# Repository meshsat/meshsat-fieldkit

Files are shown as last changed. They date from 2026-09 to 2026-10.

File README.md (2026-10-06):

# MeshSat Field Kit hardware

Hardware for the MeshSat field kits, the portable go-boxes that carry a MeshSat Bridge (a Raspberry Pi 5 in V1, three Compute Module 5 in V2) with its radios, satellite modem, cellular modem, GPS and power into the field. Since October 2026 it also holds the compact kit, the pocket-sized node (`compact/`). The software lives in the [meshsat](https://github.com/meshsat/meshsat) repository. This repository holds the mechanical and electronic design, the build records and the manufacturing files.

MeshSat is a prototype. Nothing here has been through a field deployment yet. The V1 kits are bench and demo units. The V2 boards are designed and generated, and the engineering foundations beneath them are still being completed: no V2 board is ready for layout, no layout of boards A, B, C, D, E or P carries its board's corrected schematic (E5 has none), and none has been fabricated or ordered ([`v2/docs/CURRENT-EVIDENCE.md`](v2/docs/CURRENT-EVIDENCE.md): "Foundations incomplete; 0 boards ready for layout; 0 physically verified").

## Latest: compact v2, the pocket-sized node in a printed enclosure (6 October 2026)

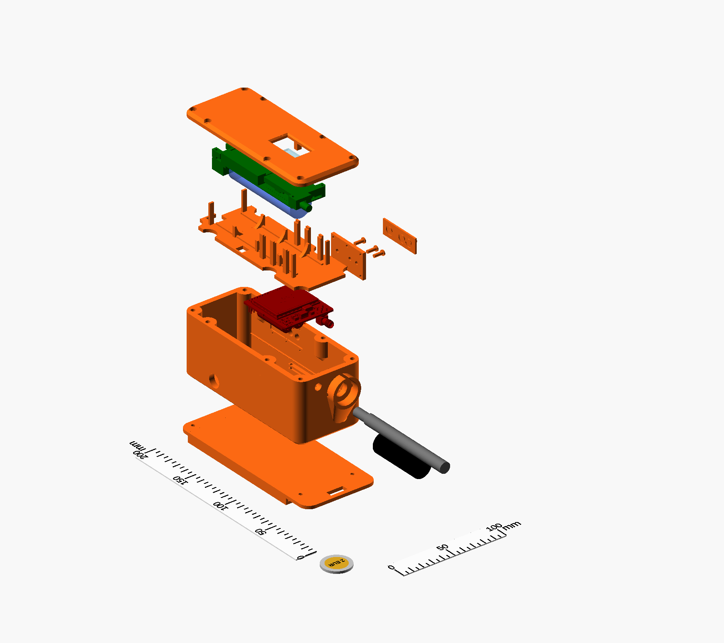
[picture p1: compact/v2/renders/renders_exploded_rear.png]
Exploded view of the compact v2 enclosure as designed: the belt plate, the body with the SOS guard and the LoRa antenna, the RockBLOCK 9704 on its rails, the separator, the T-Beam Supreme with its cell, the lid with the OLED window, and the button membrane, plungers and retainer to the side, with a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


<sub>The compact v2 enclosure exploded, as designed (an OpenSCAD render; nothing printed). From the bottom: the belt plate, the body with the SOS guard and the LoRa antenna, the RockBLOCK 9704-SMA on its rails, the printed separator, the T-Beam Supreme with its 18650 cell, the lid with the OLED window; to the side, the TPU button membrane, the three plungers and their retainer.</sub>

The compact kit is the small MeshSat node: a Meshtastic LoRa radio and an Iridium modem in a case that fits a pocket, running the MeshSat fork of the Meshtastic firmware and talking to the MeshSat phone apps over one Bluetooth link. Its third version, **compact v2**, puts a LILYGO T-Beam Supreme over a RockBLOCK 9704-SMA in a 3D-printed stacked enclosure: ASA body, lid, separator and carry plates, a TPU membrane over the board's three side buttons, an O-ring cord seal, a polycarbonate pane over the OLED, two SMA bulkheads, an IP67 panel USB-C, an M12 vent and a 12 mm IP67 switch under a guard; 62.5 x 146.0 x 62.7 mm, 154.0 mm long with the SOS guard. The design is `meshsat-enclosure` v0.6 of 5 October 2026, the answer to an engineering audit of its v0.5: both boards are registered from the makers' STEP models, every printed part is clash-checked against them, and three test coupons (the 9704 rail slot, the rim with its seal and inserts, the upper bay with the real board) come before any full print. [`compact/`](compact/README.md) holds the version table for compact v0, v1 and v2; [`compact/v2/`](compact/v2/README.md) the source, the print files, the coupons, the renders and the validation chain.

State: designed, and cleared by its own audit response for prototype printing only. The first test coupons are being printed in October 2026; nothing has been printed, fitted or sealed. Open before a full build: the panel part numbers, how the 9704 is powered, Ground Control's certification condition on other transmitters in the same housing, and the leak, button and insert tests ([`compact/v2/AUDIT-RESPONSE.md`](compact/v2/AUDIT-RESPONSE.md)). Firmware, wiring and the Bluetooth contract: [meshsat-esp32](https://github.com/meshsat/meshsat-esp32), [meshsat-firmware](https://github.com/meshsat/meshsat-firmware) and [docs.meshsat.net/node/](https://docs.meshsat.net/node/).

## News

| Date | What |
|---|---|
| 6 October 2026 | The compact kit joins this repository as [`compact/`](compact/README.md): the version table for compact v0, v1 and v2, and the v2 enclosure package (OpenSCAD source, print STLs, test coupons, renders, validation chain, the makers' reference CAD). The first test coupons are being printed. |
| 5 October 2026 | The v2 enclosure reaches v0.6, the response to an engineering audit of v0.5 (findings F01 to F15, [`compact/v2/AUDIT-RESPONSE.md`](compact/v2/AUDIT-RESPONSE.md)): boards registered from the makers' STEP models, every printed part clash-checked, grounded test coupons in place of a floating fit check, a membrane and guided plungers for the side buttons. |
| 4 October 2026 | The V2 programme adopts an execution constitution ([`v2/docs/EXECUTION-CONSTITUTION.md`](v2/docs/EXECUTION-CONSTITUTION.md)): layer deliverables with explicit dependencies, independent checking, one freeze per candidate, and separate statements of handover readiness, power-design closure and fabrication release. |
| 3 October 2026 | A panel controller firmware for board C ([`v2/firmware/panel/`](v2/firmware/panel/README.md)): a portable core with its hardware layer, a pico-sdk port and host tests. The supplier engineering-handover entry page ([`v2/docs/handover/supplier/`](v2/docs/handover/supplier/)) with a per-board BOM reader from the committed netlists. Desk work: no board exists. |
| 27 September 2026 | The case set for the Peli 1450 ([`v2/release/case-2026-09-27/`](v2/release/case-2026-09-27/README.md)): face plate, RF entry plates, connector plate, frame legs and the lid tray as CAD, drawings and 1:1 templates. Nothing cut or fitted. |
| 26 September 2026 | Circuit corrections in the schematics of boards A, B, C, D, E and P. No committed layout carries them; the deliverable folders of `v2/release/revA/` predate them. |
| 7 September 2026 | The MESHSAT-830 generation: the Peli 1450 go-box around three Compute Module 5 slots, its boards generated from their generators (the V2 section below). |
| 3 September 2026 | This repository opens with the Rev A design release (`revA`) of the previous board generation (one compute module, the Touch Display, a twelve-cell battery module), kept on the GitHub release as the record. |
| April 2026 | The V1 kits tesseract and parallax built, in use since as bench and demo units ([`v1/`](v1/README.md)). |

## Folders

| Folder | What it is | State |
|---|---|---|
| `v1/` | tesseract and parallax as built: IP67 case, HDPE plates on M3 rods, UV-K5 + AIOC APRS chain, per-kit BOM and GPIO pinouts, FreeCAD plate model | built April 2026, in use |
| `v2/` | the Peli 1450 go-box of the MESHSAT-830 generation: seven carrier PCBs around three Compute Module 5 slots, an aluminium control face on the 1450PF panel frame with a sealed monitor in it and a backer board under it, a removable stack on a floor dock, a 4S pack built for the kit (about 145 Wh) in the east pocket | first generated 7 September 2026; circuits corrected on 26 September 2026 in the schematics only; foundations incomplete, 0 boards ready for layout, nothing built or ordered |
| `compact/` | the compact kit, the pocket-sized node: the version table for v0 (XIAO ESP32-S3 + Wio-SX1262 + RockBLOCK 9603 bench unit), v1 (LILYGO T-Beam Supreme + RockBLOCK 9603 for a Peli 1020) and v2 (T-Beam Supreme over a RockBLOCK 9704-SMA in a 3D-printed stacked enclosure, OpenSCAD, in `compact/v2/`) | v0 and v1 are bench units running since September 2026 (the v1 Peli build is not finished); v2 designed 5 October 2026, cleared by its own audit response for prototype printing only, nothing printed or fitted |

## V1: tesseract and parallax

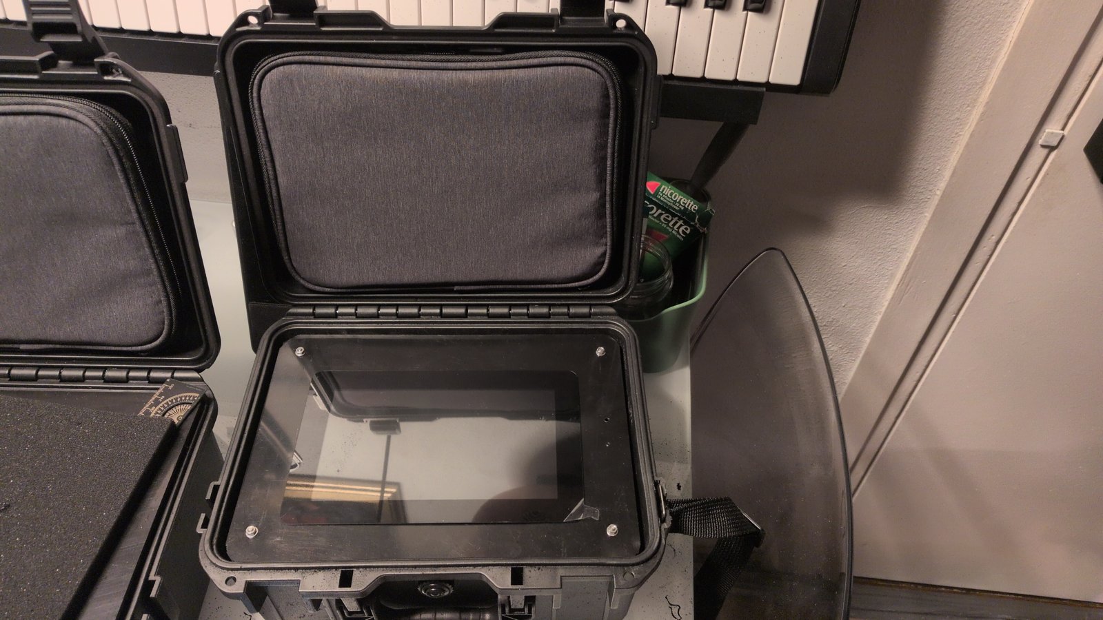
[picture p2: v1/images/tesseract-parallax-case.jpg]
tesseract, one of the two V1 kits, in its IP67 case with the display under the top plate


Two hand-built kits that differ only in the satellite modem (tesseract: RockBLOCK 9603 SBD, parallax: RockBLOCK 9704 IMT). Pi 5 with a Geekworm X1202 UPS, LilyGO T-Call A7670E, u-blox GPS, Quansheng UV-K5(8) with an AIOC for APRS, ESP32-S3 LoRa for Meshtastic, RTL-SDR v4, ZigBee CC2652P, DCF77 receiver, WeAct 3.7 inch e-paper, Raspberry Pi Touch Display 2, all on three HDPE plates in an IP67 case with SMA bulkheads. Details, BOM and pinouts in [`v1/README.md`](v1/README.md). **To build one: [`v1/BUILD.md`](v1/BUILD.md)** (parts, case drilling, plates, harness tables, software provisioning, checks).

## V2: the carrier set (MESHSAT-830 generation, 7 September 2026)

Seven KiCad 9 boards replace the plates, the loose wiring and the USB hub. Three Raspberry Pi Compute Module 5 sit in identical slots on one carrier, each with a PCIe switch, an NVMe drive, a USB 3 hub and a card slot; most radios and the sensor and panel controllers are USB devices on those hubs, shared by the HAL across the three modules, which run k3s; each of the three hub banks is designed to switch in hardware from its home module to a neighbour, decided by three I/O supervisors voting two of three, so losing a module is meant to move its USB peripherals instead of removing them. Not everything is on a hub: the two WiFi link cards are PCIe cards on two different modules, and only their antennas move; the compute modules' own WiFi and Bluetooth stay with each module; and two bearers have no second path and go with their module, the LoRa module on one module's SPI and the 5G data path on another's PCIe lane ([`v2/docs/ARCH-PCB-B-IOHA.md`](v2/docs/ARCH-PCB-B-IOHA.md) section 15). The stack (PCB-A power with the VHF mezzanine, PCB-B compute) lifts straight out of the case, and a dock strip on the case floor carries the 9 to 36 V front end, the solar tracker, the sensor controller and the contact block that the stack lands on; as generated, eleven antenna paths blind-mate at the same time (a twelfth, the third 5G jack, waits on the board E clamp fit under owner ruling D-07). The face is a 3 mm aluminium plate on the Peli 1450PF frame (over Peli's o-ring, case choice C1) with a Xenarc IP67 monitor set into it, a wide-temperature e-paper under a lens, sealed switches, two headset jacks and a camera window, with the backer board C7 (an RP2040 panel controller) under it and the 30 W VHF amplifier bolted to its underside. The pack is a 4S lithium-ion pack, built rather than bought, for the pocket beside A24 at the east wall (the BB-2590/U did not fit the case; appendix 32.62). On 26 September 2026 the owner ruled its size: one 4S3P block of Samsung INR18650-35E cells, about 145 Wh, shrink-wrapped in that pocket, its fit designed against Peli's own figures ([`v2/docs/CASE-MARGINS.md`](v2/docs/CASE-MARGINS.md)), with missions longer than the pack relying on vehicle or solar input. The product brief, the concept of operations with its PROVISIONAL runtime per power state, the device set and the qualification plan are in [`v2/docs/PRODUCT-BRIEF.md`](v2/docs/PRODUCT-BRIEF.md), [`v2/docs/CONOPS.md`](v2/docs/CONOPS.md), [`v2/docs/V2-SPEC.md`](v2/docs/V2-SPEC.md) and [`v2/docs/TEST-PLAN.md`](v2/docs/TEST-PLAN.md); none of it has been built. Against Peli's own figures, the antenna entries are twelve gas-discharge arrestors on one RF entry plate per end wall at 59 mm and the wall items share one connector plate between the hinge fairings, choices the design session took under the owner's standing rule of 26 September 2026 ([`v2/docs/CASE-MARGINS.md`](v2/docs/CASE-MARGINS.md) section 4); the case generators carry them since `c351115d` and the current case set, CAD, drawings and 1:1 templates, is [`v2/release/case-2026-09-27/`](v2/release/case-2026-09-27/README.md), while the committed board files and the deliverable folders of `v2/release/revA/` predate it.

| Board | Rev (newest deliverable folder) | Declared phase | Size (mm) | Layers | Role |
|---|---|---|---|---|---|
| PCB-A POWER + I/O | A24 | A32 | 240 x 160 | 6 | the 14.4 V node from the 4S pack, BQ25731 SMBus charger, three 5.1 V slot rails and a device rail, the 13.8 V amplifier rail and the 12 V HF rail (both EMCON gated), the 54 V PoE rail, the 45 W USB-C outlet, INA226 rail monitors, the D8 mezzanine site, eleven blind-mate RF receptacles, the dock contacts |
| PCB-B COMPUTE | B19 (quote only, not routed) | B21 | 330 x 200 | 6 (an 8-layer trial ruled 25 Sep 2026) | three Compute Module 5 slots on board-to-board receptacles, per slot a PCIe switch with an NVMe 2242 and a card slot (a WiFi link card, the 5G module, the second WiFi link card), a four-port USB 3 hub and a cooler fan; the KSZ9897 Ethernet switch to the wall port with PoE, the three-input HDMI switch to the monitor, the LimeSDR bay, the RockBLOCK site, the LG290P GNSS, the E22 1 W LoRa module, two E72 radios (Zigbee and Thread), the holdover clock, the secure element, the panel ribbon |
| PCB-C PANEL BACKER | C24 | C24 | 344 x 228 ring | 4 (6 ruled 25 Sep 2026, not yet regenerated) | the ring under the face plate: the RP2040 panel controller (a USB device with the hardware EMCON and ZEROIZE lines), the sixteen LEDs under IP68 light guides (and, in the schematic since its round 8, a seventeenth, the hardware EMCON lamp, whose light guide in the plate is owed), two GPIO expanders, the e-paper flex socket and its boost stage, the sounder driver, the ambient light sensor, the lands for the sealed switches, the holes for the headset jacks and the monitor's connector block |
| PCB-D VHF APRS | D11 | D12 | 100 x 80 | 4 | the NiceRF SA868 exciter, the T/R relay, the low-pass filter and the leads to the RA30H1317M1 30 W module on the plate, a USB audio codec and headphone amplifier for the two headset jacks, a USB hub and the control bridge, the PTT and EMCON logic, the amplifier gate bias switch |
| PCB-E1 DOCK STRIP | E9 | E17 | 267 x 68 | 4 | the floor strip: 9 to 36 V vehicle and shore entry with the LM5176 front end, the solar tracker, the pack entry with its fuse and SMBus, the sensor controller (a second RP2040) with the climate, seal, water, gas, motion, lightning, Geiger and outside-pod inputs, two mixer fans, one blind-mate clamp bar with twelve cavities (board A's eleven RF sites and the third 5G jack of owner ruling D-07), the raised contact block |
| PCB-E5 DOCK BLOCK | E5 | E5 (no schematic) | 43 x 26 | 2 | the raised block on the strip: the targets the stack's spring pins land on, wire lands underneath |
| PCB-P PACK BMS | P4 | P4 | 70 x 44 | 2 (4 at 2 oz ruled 25 Sep 2026, not yet regenerated) | inside the 4S pack: the BQ4050 SMBus gauge with protection and balancing, two high-side N-FETs, the 2 mohm shunt, the 25 A blade, the cell tap, thermistor and SMBus headers, the lead lands (appendix 32.62) |

The revision column names the newest deliverable folder in `v2/release/revA/boards/`, and the declared phase is the board this project is building ([`v2/docs/CURRENT-EVIDENCE.md`](v2/docs/CURRENT-EVIDENCE.md)). Every deliverable folder predates the circuit corrections of 26 September 2026 (`faf8c981`, `458b2873`, `d90f30e4`) and every later one, which are in the schematics only: no layout of boards A, B, C, D, E or P carries its board's corrected netlist (E5 has no schematic). The renders below show those older layouts.

**Reading this page inside an engineering handover snapshot** (`v2/release/handover/<version>.zip`): the snapshot leaves out `v2/images/` (renders, presentation) and `v1/` (the V1 kits, out of the V2 handover's scope), so the images below and the links into `v1/` do not resolve there; they do in this repository. The snapshot's `EXCLUDED.tsv` lists every file left out, and its `START-HERE.md` section 7 says why.

| | |
|---|---|
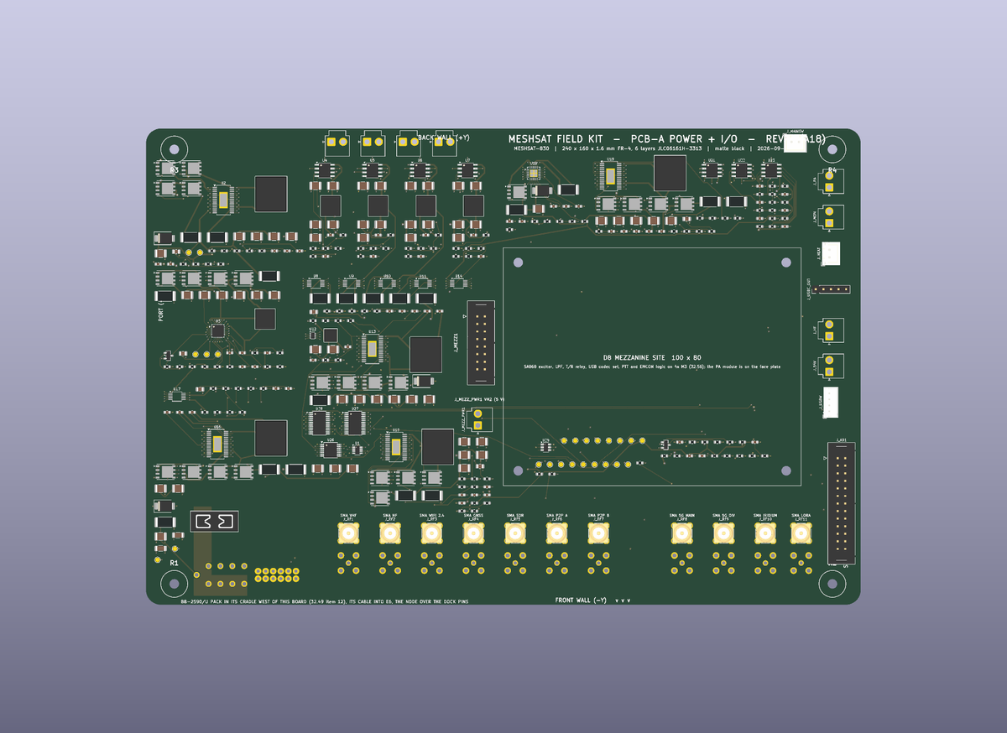
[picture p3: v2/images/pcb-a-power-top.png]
PCB-A
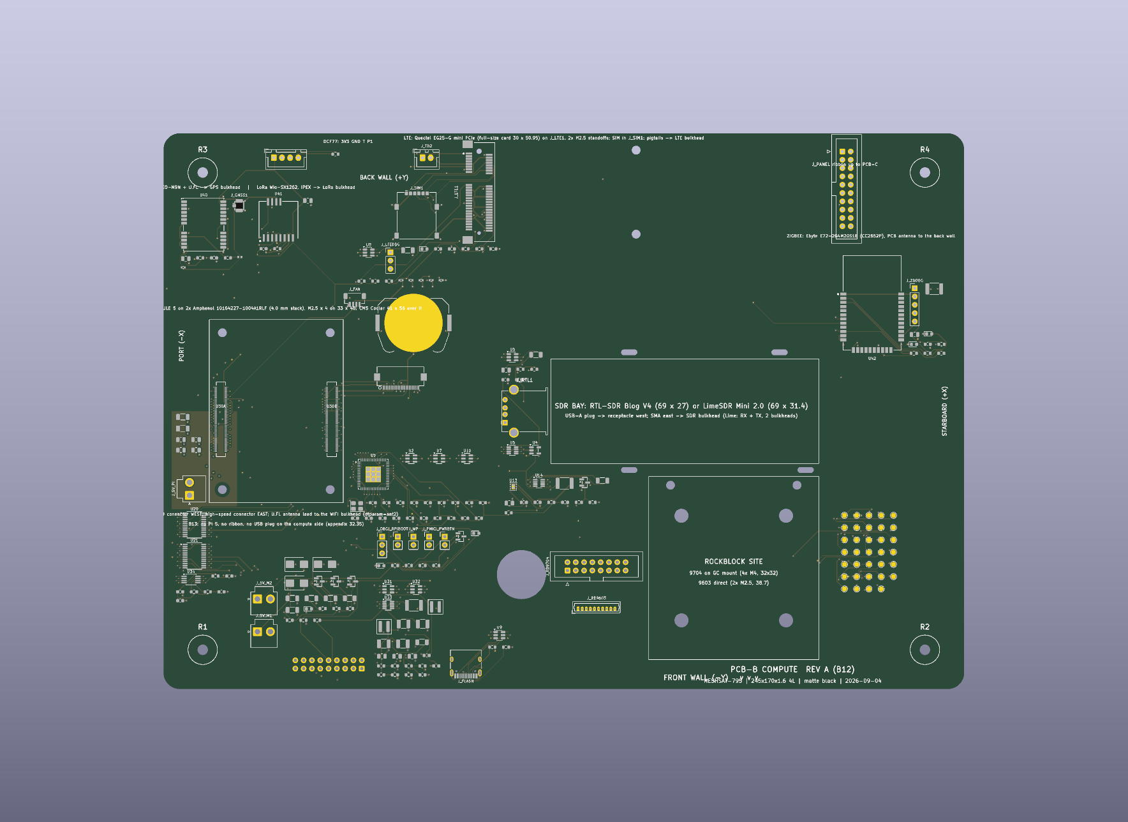
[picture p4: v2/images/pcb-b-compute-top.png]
PCB-B
|  |  |
| PCB-A POWER + I/O | PCB-B COMPUTE |
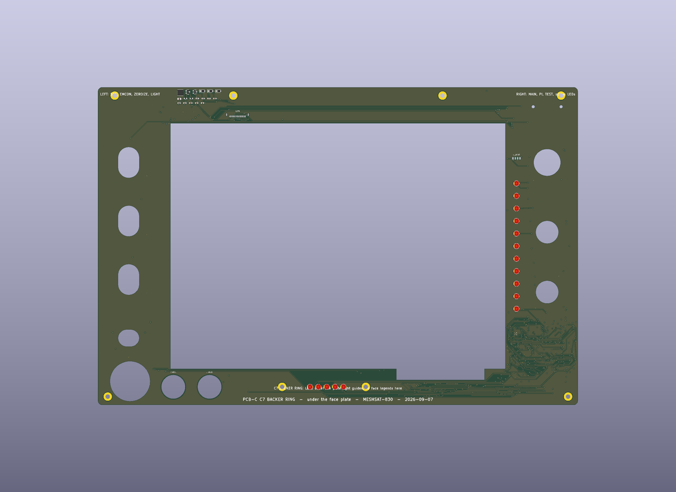
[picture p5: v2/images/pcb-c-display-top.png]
PCB-C
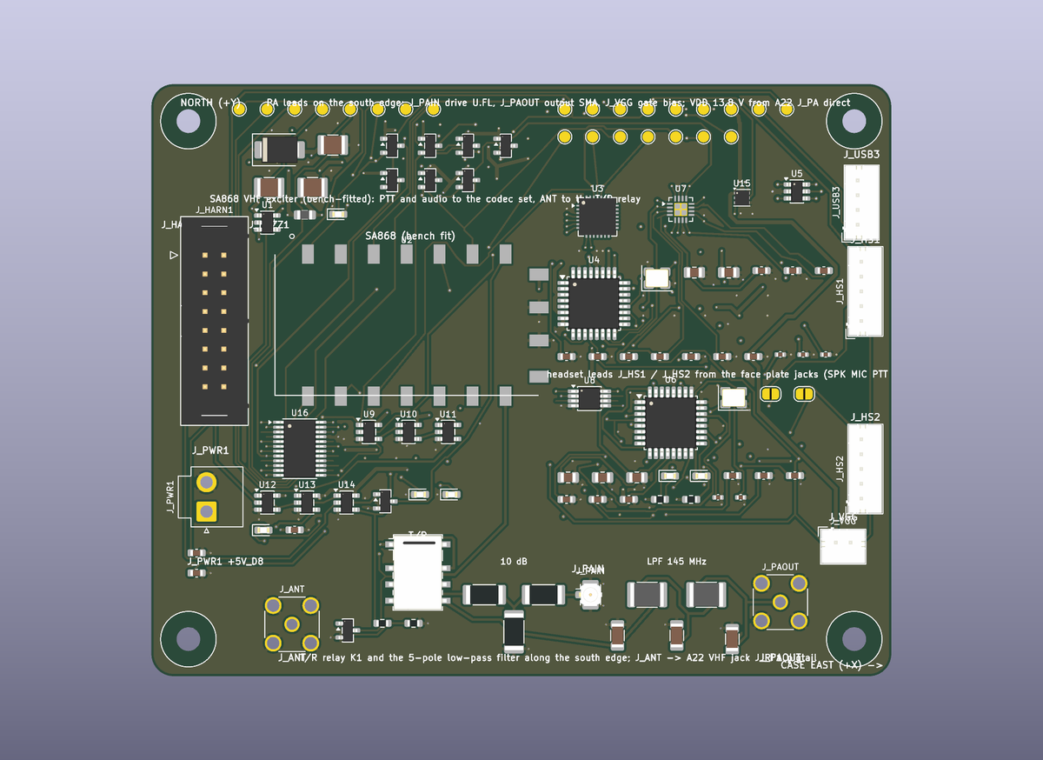
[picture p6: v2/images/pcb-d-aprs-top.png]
PCB-D
|  |  |
| PCB-C PANEL BACKER | PCB-D VHF APRS |
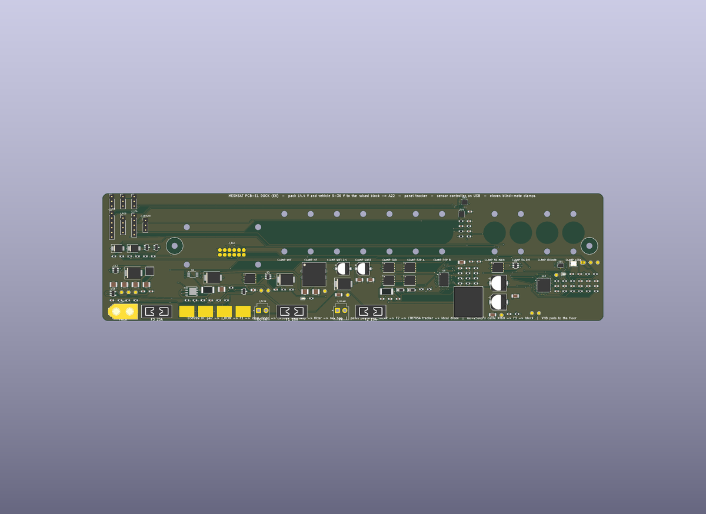
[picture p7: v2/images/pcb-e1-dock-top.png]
PCB-E1
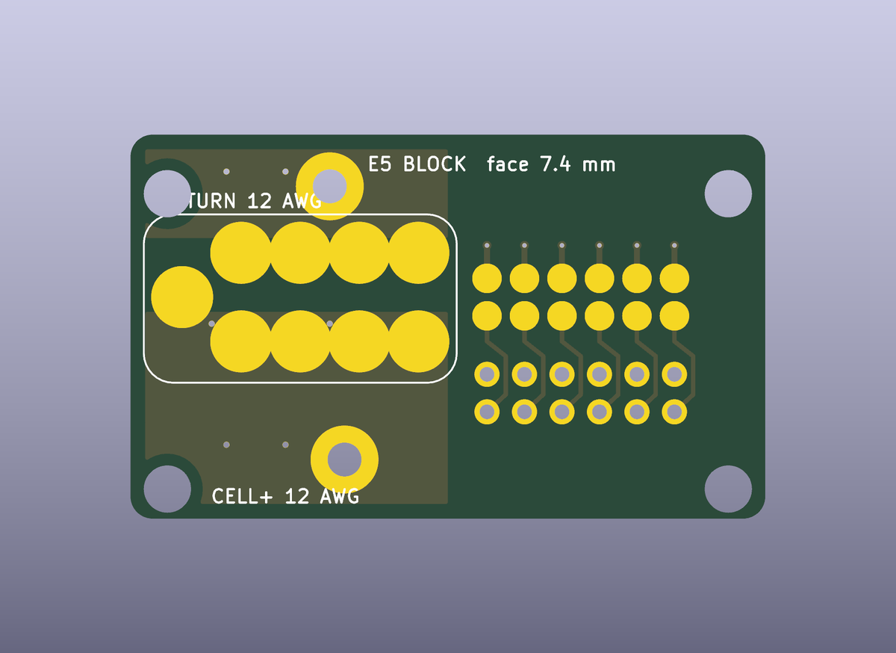
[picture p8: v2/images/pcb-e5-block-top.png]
PCB-E5
|  |  |
| PCB-E1 DOCK STRIP | PCB-E5 DOCK BLOCK |
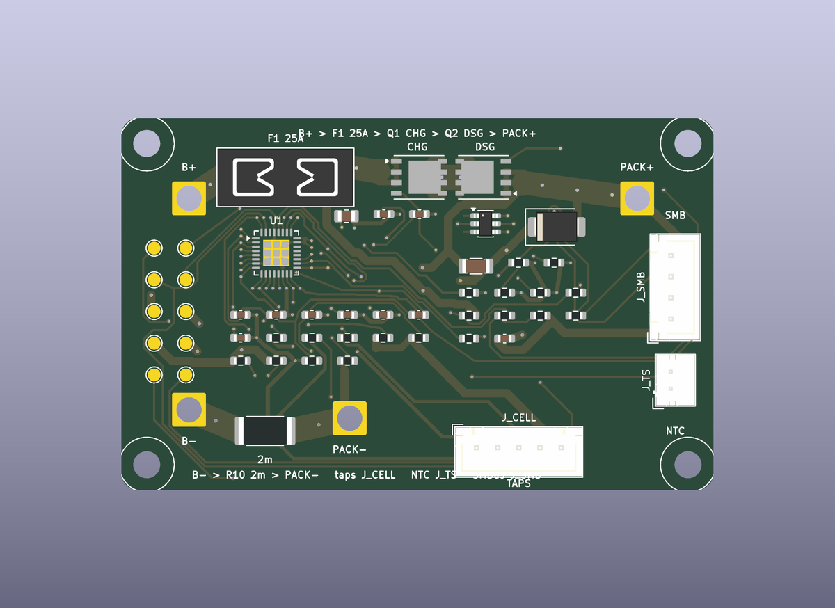
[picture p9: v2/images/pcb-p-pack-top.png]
PCB-P
|  | |
| PCB-P PACK BMS | |

Concept renders of the assembled kit as designed (not built; `v2/cad/render/` holds the Blender scene, `v2/images/concept-1450/README.md` the full set):

| | |
|---|---|
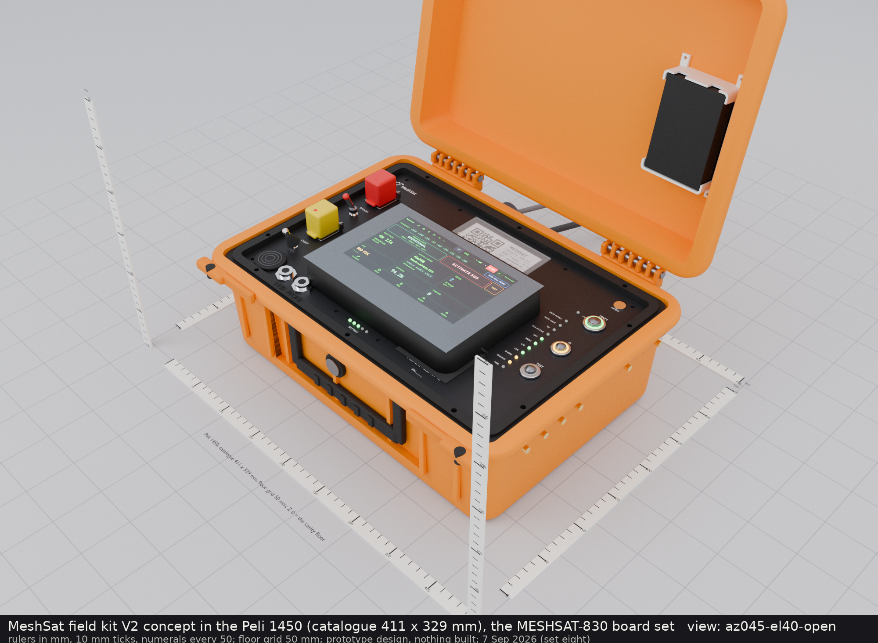
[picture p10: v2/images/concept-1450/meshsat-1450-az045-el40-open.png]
overview
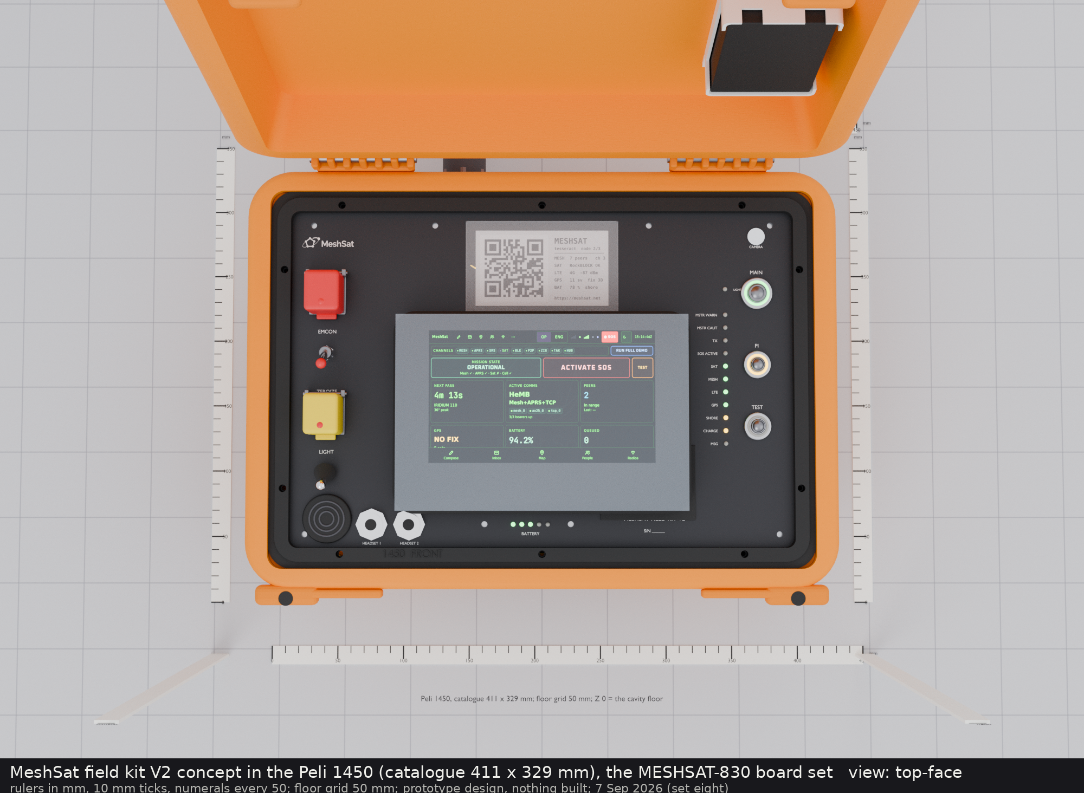
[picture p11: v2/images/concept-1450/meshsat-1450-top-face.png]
face
|  |  |
| the open case from the front | the face from above |
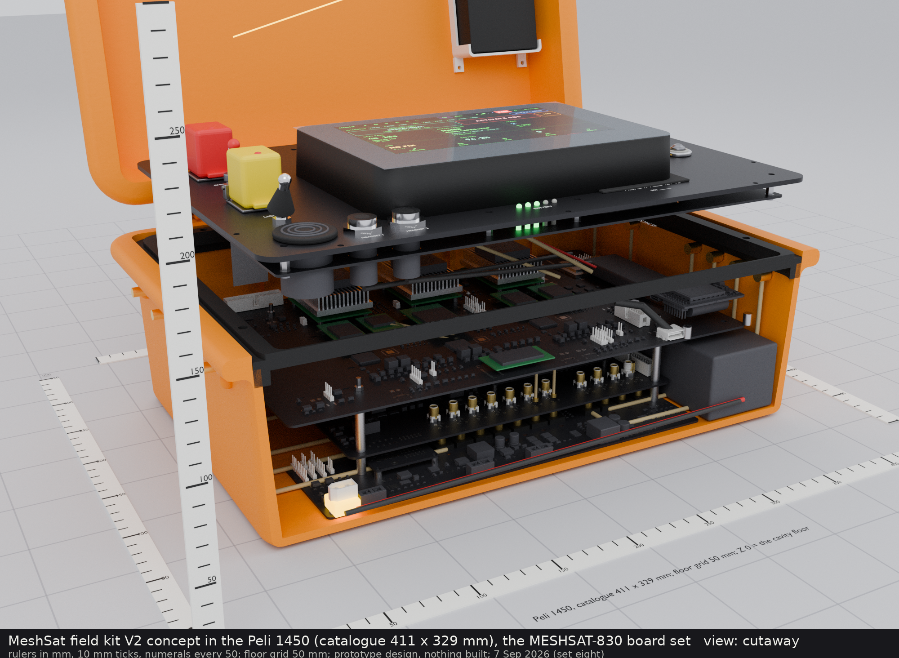
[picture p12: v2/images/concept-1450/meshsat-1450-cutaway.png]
cutaway
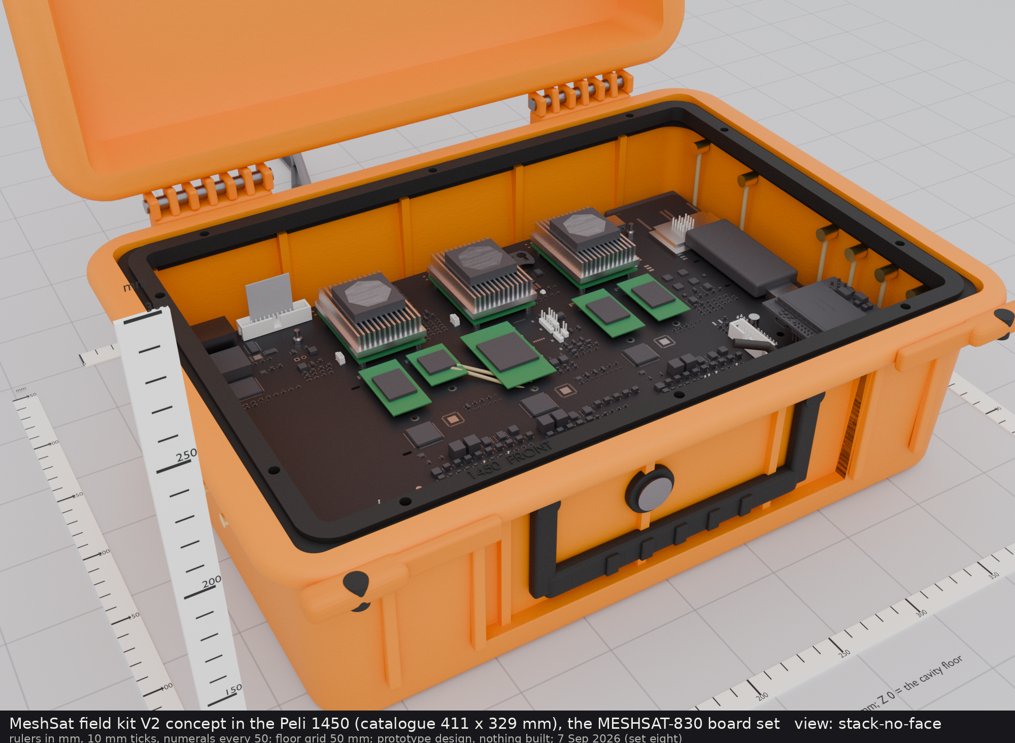
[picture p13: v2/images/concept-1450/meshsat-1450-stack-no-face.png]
stack
|  |  |
| the front wall cut away and the face lifted | the stack without the face |
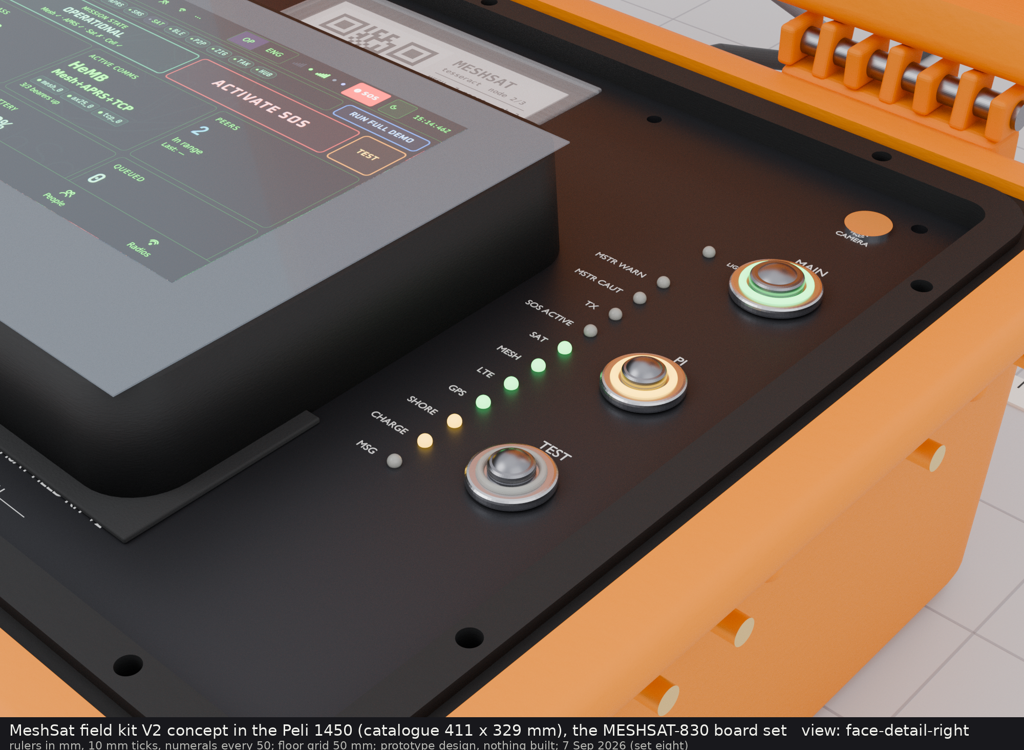
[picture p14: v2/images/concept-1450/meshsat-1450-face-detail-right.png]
detail
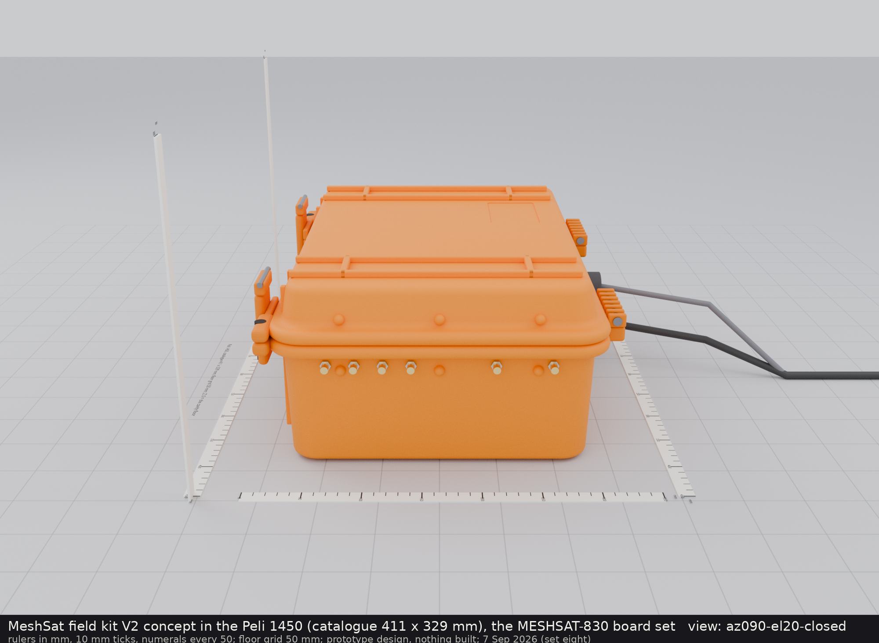
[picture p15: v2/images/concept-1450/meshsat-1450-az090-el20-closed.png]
closed
|  |  |
| the switch corner | closed for transport |

**The V2 build guide, [`v2/BUILD.md`](v2/BUILD.md), is the 7 September generation's guide, kept as the assembly narrative and not to be used to order boards:** no board is ready for layout, and the order folder is rebuilt and quarantined with nothing ordered from it (owner decision 41 of 25 September 2026). Sources, generators, vendor references, the release and the order record are described in [`v2/README.md`](v2/README.md). The design record is [`v2/docs/MESHSAT-709-geometry-appendix.md`](v2/docs/MESHSAT-709-geometry-appendix.md), the build procedure [`v2/docs/ASSEMBLY.md`](v2/docs/ASSEMBLY.md), the panel controller contract [`v2/docs/PANEL.md`](v2/docs/PANEL.md).

## How to build one

| | Guide | What it covers |
|---|---|---|
| V1 | [`v1/BUILD.md`](v1/BUILD.md) | the 33-line parts list per kit, bulkhead and hole schedule, the three HDPE plates and the rod stack, what goes on which floor, the GPIO harness tables for both kits as wired, the Pi 5 provisioning sequence and its traps, the checks that prove the kit works |
| V2 | [`v2/BUILD.md`](v2/BUILD.md) | the 7 September generation's guide, headed as history and not for ordering (decision 41; 0 boards ready for layout): the boards as generated, everything else to buy, case and frame preparation, the 4S pack, the assembly order with torques, leads and pigtails, coating and labels, software bring-up, the open items, with the lines that contradict the current baseline corrected in place |

## Working with this repository

- Binaries (STEP, FreeCAD, DXF, zips, PDFs, renders) are ordinary git objects; a clone is about 400 MB and needs no Git LFS.
- KiCad 9, Freerouting and the generator scripts run headless on a rented build host; see `v2/README.md` for the pipeline and the prerequisites.
- `v2/vendor/` holds third-party reference material (manufacturer CAD, datasheets) under the vendors' own terms; see `v2/vendor/README.md`.

## Licence

The hardware design, documentation and generator scripts in this repository are released under the CERN Open Hardware Licence Version 2, Strongly Reciprocal (CERN-OHL-S-2.0), see [`LICENSE`](LICENSE). Third-party files under `v2/vendor/` are not covered by it.

## Links

- Project site: [meshsat.net](https://meshsat.net)
- Bridge software: [github.com/meshsat/meshsat](https://github.com/meshsat/meshsat)
- This repository on GitHub: [github.com/meshsat/meshsat-fieldkit](https://github.com/meshsat/meshsat-fieldkit) (mirror of the GitLab original)

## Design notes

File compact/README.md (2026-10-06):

# Compact kit: the pocket-sized MeshSat node

The compact kit is the small MeshSat node: a Meshtastic LoRa radio and an Iridium modem in a case that fits a pocket, running the MeshSat fork of the Meshtastic firmware and talking to the MeshSat phone apps over one Bluetooth link. It is a kit in its own right beside the field kits of `v1/` and `v2/`, with its own version line. This folder holds the hardware side: the version table below and, under `compact/v2/`, the enclosure design. The firmware, the wiring tables, the bench tools and the Bluetooth contract live in [meshsat-esp32](https://github.com/meshsat/meshsat-esp32) and [meshsat-firmware](https://github.com/meshsat/meshsat-firmware); the user guide is [docs.meshsat.net/node/](https://docs.meshsat.net/node/).

MeshSat is a prototype. The v0 and v1 nodes are bench units. The v2 enclosure is a design: nothing of it has been printed or fitted, and its own audit response clears it for prototype printing only.

## Versions

| | v0 (bench) | v1 (prototype) | v2 (design) |
|---|---|---|---|
| Board | Seeed Studio XIAO ESP32-S3 + Wio-SX1262 | LILYGO T-Beam Supreme (ESP32-S3, SX1262, u-blox M10S GPS) | LILYGO T-Beam Supreme |
| Satellite | RockBLOCK 9603 (Iridium SBD) | RockBLOCK 9603 (Iridium SBD) | RockBLOCK 9704-SMA (Iridium IMT) with Ground Control's helical antenna |
| Power | USB power bank | one 18650 cell in the T-Beam's holder, charged over USB-C; the modem runs from the T-Beam's power chip | one 18650 cell in the T-Beam's holder; how the 9704 is fed is an open item of the design (Ground Control's battery window for it is 3.6 to 4.5 V) |
| Case | Peli 1050 | Peli 1020 with an IP68 USB-C port and a panel power button; the build is not finished | a 3D-printed stacked enclosure: the 9704 on edge rails in the lower bay, a printed separator, the T-Beam and its cell in the upper bay, an OLED window in the lid; ASA parts, a TPU button membrane, an O-ring cord seal, a polycarbonate pane, two SMA bulkheads, an IP67 panel USB-C, an M12 vent, a 12 mm IP67 switch, a MOLLE or belt plate; 62.5 x 146.0 x 62.7 mm, 154.0 mm long with the SOS guard |
| Firmware env | `meshsat-xiao-s3-rockblock` | `meshsat-tbeam-s3-rockblock` | not part of this package: firmware and app support for the 9704 on the node is not claimed here |
| State | tested on the bench, September 2026; retired from the phone role on 21 September 2026 | running since 21 September 2026 on the bench and in a garden | designed 5 October 2026 (`meshsat-enclosure` v0.6); the first test coupons are being printed in October 2026; nothing printed or fitted |

The v0 and v1 wiring (four wires between the board and the RockBLOCK) and the proven table are in the meshsat-esp32 README and on docs.meshsat.net/node/build; they are not repeated here.

## v2: the printed enclosure (`compact/v2/`)

`compact/v2/` is the OpenSCAD package `meshsat-enclosure-v0.6` as delivered on 5 October 2026, the design's response to an engineering audit of its v0.5 (findings F01 to F15, each answered in [`v2/AUDIT-RESPONSE.md`](v2/AUDIT-RESPONSE.md)). Its own [`README.md`](v2/README.md) is the print and assembly guide: the print order (three test coupons first, then one full prototype in PLA or PETG, then the ASA set), materials and orientations, the hardware list, the assembly notes and the electrical items it leaves open.

| Path | Content |
|---|---|
| `v2/source/meshsat-enclosure-v0.6.scad` | the design, one file; `PART` selects a printable part, a coupon, the assembly or the exploded view |
| `v2/print-stl/` | the eight printable parts, exported in print orientation: body, lid, separator, membrane (TPU), plungers (three), retainer, MOLLE plate, belt plate |
| `v2/coupons/` | the three test coupons: `rails` (the 9704 slot fit), `rimlid` (seal groove, inserts, lid screws), `board` (the upper bay with the separator, the real T-Beam and the lid) |
| `v2/renders/` | assembly, two exploded views (with a ruler and a 2 EUR coin) and the button detail |
| `v2/validation/` | `build_and_check.sh` regenerates every STL and reruns the checks; `clash_check.py` intersects every printed part, in assembled position, with the makers' board geometry; `mesh_report.py` writes the printability report with a SHA-256 per STL; `build/` holds the results for this release (clash 0.000 mm3 against both boards, the self-checks as expected) |
| `v2/reference-cad/` | the makers' models the boards were registered from (LilyGO, Ground Control), with their own [`README.md`](v2/reference-cad/README.md): not covered by this repository's licence |

Two files of the delivered package are not duplicated here because this repository already holds them byte for byte: the RockBLOCK 9704-SMA board STEP (`v2/vendor/rockblock/RockBLOCK 9704-SMA-2A.step`, 52.7 MB) and the mount drawing (`v2/vendor/rockblock/rb9704-sma-dims.pdf`). The validation chain reads only the tessellated meshes in `v2/reference-cad/meshes/`, so it runs without them. The package as delivered: `meshsat-enclosure-v0.6.zip`, 58 files, sha256 `002b31a9390fab535e158f40d89099b727800e5863262c885cb629dfd9aa1761`. Its README and audit response are kept as delivered, with their dashes written out under this repository's drafting rule (ranges as "a to b", empty evidence cells as "none"); nothing else in them changed.

Open before a full build, in the design's own words (the matrix in `v2/AUDIT-RESPONSE.md`): the exact panel part numbers and their cut-outs (F11); how the 9704 is powered (F12); Ground Control's certification condition that no other transmitter sits in the same housing as the 9704, where this design puts LoRa, Bluetooth and WiFi beside it (F13, their written position is owed); the leak, button and insert tests and the qualification sequence (F14); and the real-part fit of the 1.80 mm rail slot and of the 18650 holder, which is not in LilyGO's STEP. The next revision, v0.7, is owed before the full set is printed: a flip cover over the SOS button and the final panel hardware.

## Licence

The enclosure design (the `.scad` source and the STL files made from it) is released under this repository's licence, CERN-OHL-S-2.0. The files under `v2/reference-cad/` belong to their makers and are reference material only; see that folder's README.

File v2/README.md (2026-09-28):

# V2: the Peli 1450 carrier set (MESHSAT-830 generation)

Seven KiCad 9 boards for the kit V2 go-box: a Peli 1450 case with the 1450PF panel frame. The power and compute boards stack on four M3 rods and lift out of the case in one piece; a dock strip on the case floor carries the 9 to 36 V front end, the solar tracker, the sensor controller and the raised contact block that the stack blind-mates onto, with eleven antenna paths mating at the same time as generated (twelve with the third 5G jack of owner ruling D-07, which waits on the board E clamp fit). The control face is a 3 mm aluminium plate on top of the frame, over Peli's o-ring and screwed into Peli's inserts (`cad/face_plate.py`, `release/case-2026-09-27/face-plate/`; the session's case choice C1 of `docs/CASE-MARGINS.md` section 4, which the case generators carry since `c351115d`) with a Xenarc 709GNK monitor set into it, its glass level with the aluminium face (owner ruling of 9 September 2026, appendix 32.85), the backer board C7 hanging under it and the 30 W VHF module bolted to its underside; the 4S pack, built for the kit rather than bought (one 4S3P block of about 145 Wh by the owner's ruling of 26 September 2026, its fit designed against Peli's own figures, `docs/CASE-MARGINS.md`), lies in the pocket at the east end wall (appendix 32.62), and the antenna entries are twelve gas-discharge arrestors on one RF entry plate per end wall at 59 mm (case choices C2 and C4, carried by the case generators and the case set `release/case-2026-09-27/` since `c351115d`; the committed board files and the deliverable folders of `release/revA/` predate them). Nothing here has been built: the boards are designed and generated, no board is ready for layout (`docs/CURRENT-EVIDENCE.md`: "Foundations incomplete; 0 boards ready for layout; 0 physically verified"), and no set has been ordered.

The rulings that bind the design (details in `docs/MESHSAT-709-geometry-appendix.md`, sections 32.49 to 32.61, and the specification `docs/V2-SPEC.md`): three identical Compute Module 5 slots with most radios and the sensor and panel controllers USB devices shared by the HAL, k3s across the modules, and each hub bank switchable in hardware between its home module and a neighbour so one module's loss is meant to move its USB peripherals rather than remove them; the two WiFi link cards are PCIe cards on two modules whose antennas, not the cards, move, the compute modules' own radios stay with each module, and the LoRa module (one module's SPI) and the 5G data path (another's PCIe lane) have no second path and go with their module (`docs/ARCH-PCB-B-IOHA.md` section 15); the pack, the charger and the power control on PCB-A; no vent opening anywhere in the case; EMCON a hardware line from the panel toggle, plus a software hold, meant to silence every transmitter, with the radios dark and only the VHF receiver, GNSS, DCF77 and the lightning sensor still listening (the owner's ruling of 26 September 2026): as generated at `45bde541` it is drawn to remove the supply of the SDR, the RockBLOCK, the LoRa module, both Zigbee and Thread radios, the HF unit and both WiFi link cards, to turn off the amplifier's rail and keying while the VHF exciter keeps receiving, to pull the compute modules' own WiFi and Bluetooth disables low, and to put the 5G module in airplane mode through its disable pin, and since board B's round 8 (27 September 2026) it also removes the 5G module's supply by hardware at once (SD-EMC-1r8; `docs/CONOPS.md` section 4b, `docs/feasibility/EMCON.md` section 4b); read transmitter by transmitter (`docs/feasibility/EMCON.md` section 0a) none of the kit's 17 transmitters is dark end to end: the radio's own chain closes at desk for 15 and is open for the SA868 (its PTT pin's receive threshold is unpublished) and the RockBLOCK 9704 (once its supply is cut it runs on its own supercapacitors with its ENABLE held by firmware, so the ENABLE forced low by the EMCON hardware is owed); every row also waits on the items the rows share (the toggle and its conductor, whose hardware EMCON lamp is drawn on board C since its round 8 with its light guide in the plate owed) and on the latency the session set (1 s, 20 s for a running 5G module; REQ-071), and no row has been shown on a bench (feasibility blocker FEA-002); the panel a USB device driven per `docs/PANEL.md`.

| Board | Rev (newest deliverable folder) | Declared phase | Size (mm) | Layers | Project | Deliverable folder |
|---|---|---|---|---|---|---|
| PCB-A POWER + I/O | A24 | A32 | 240 x 160 | 6 | `ecad/pcb-a-power-a23/` | `release/revA/boards/meshsat-pcb-a-revA-A24/` |
| PCB-B COMPUTE | B19 | B21 | 330 x 200 | 6 (8-layer trial ruled 25 Sep 2026) | `ecad/pcb-b-compute-b19/` | `release/revA/boards/meshsat-pcb-b-revA-B19-quote/` (quote only: placed, not routed) |
| PCB-C PANEL BACKER | C24 | C24 | 344 x 228 ring | 4 (6 ruled 25 Sep 2026, not yet regenerated) | `ecad/pcb-c-display-c8/` | `release/revA/boards/meshsat-pcb-c-revA-C24/` |
| PCB-D VHF APRS | D11 | D12 | 100 x 80 | 4 | `ecad/pcb-d-aprs-d9/` | `release/revA/boards/meshsat-pcb-d-revA-D11/` |
| PCB-E1 DOCK STRIP | E9 | E17 | 267 x 68 | 4 | `ecad/pcb-e1-dock-e7/` | `release/revA/boards/meshsat-pcb-e-revA-E9/` |
| PCB-E5 DOCK BLOCK | E5 | E5 (no schematic) | 43 x 26 | 2 | `ecad/pcb-e5-block/` | `release/revA/boards/meshsat-pcb-e5-revA-E5/` |
| PCB-P PACK BMS | P4 | P4 | 70 x 44 | 2 (2 oz; 4 at 2 oz ruled 25 Sep 2026, not yet regenerated) | `ecad/pcb-p-pack-p2/` | `release/revA/boards/meshsat-pcb-p-revA-P4/` |

Every deliverable folder in this table predates the circuit corrections of 26 September 2026 (`faf8c981`, `458b2873`, `d90f30e4`) and every later one, which are in the schematics only: no layout of boards A, B, C, D, E or P carries its board's corrected netlist (SCH-002 reads FAIL on A and B and INCONCLUSIVE on C, D, E and P; E5 has no schematic, and its board file is its design), and each board's remaining layout-entry blockers are listed in `docs/CURRENT-EVIDENCE.md`.

The previous generation (A21, B15, C6, D7, E4, E5 with a single Compute Module, the Touch Display and a twelve-cell battery module) stays on the `revA` GitHub release and in the git history as the record; its deliverable folders are replaced as the new boards land.

**Build guide: [`BUILD.md`](BUILD.md)** is the 7 September generation's guide, kept as the assembly narrative and headed as not for ordering (owner decision 41; no board is ready for layout). This page is the map of the folder.

## Layout

| Path | Content |
|---|---|
| `docs/` | `MESHSAT-709-geometry-appendix.md` (the design record, every number and every ruling), `ASSEMBLY.md` (fasteners, torque, coating, removal procedure, bench-fit lists), `PANEL.md` (the software contract for the control panel, MESHSAT-773), `V2-SPEC.md` (the approved specification of the next generation, MESHSAT-830, with its corrections of 26 September 2026), `TEST-PLAN.md` (its qualification plan), `PRODUCT-BRIEF.md` and `CONOPS.md` (the product brief and the concept of operations of the foundation baseline, MESHSAT-1357), `CURRENT-EVIDENCE.md` (what each board's evidence shows today), `CASE-MARGINS.md` (the case held against Peli's own figures, with the case choices C1 to C6), `ARCHITECTURE.md` and `feasibility/` (the architecture and the feasibility of the core functions), `EXECUTION-PLAN.md` (the foundation programme and its stage gates), `records/` (the session records the pages cite) and `reviews/` (the owner's reviews and prompts) |
| `ecad/` | the KiCad sources: one project folder per board, `meshsat.pretty/` (project footprints), `tools/` (the generators and the pipeline scripts) |
| `vendor/` | third-party reference CAD and datasheets (see `vendor/README.md`) |
| `release/revA/boards/` | the Rev A deliverables: KiCad project snapshot, Gerber zip, BOM, CPL, DRC report, schematic PDF, renders, 1:1 print |
| `release/revA/order/` | the JLCPCB order set: per-board upload folder with `ORDER-NOTES.txt`, `ORDER-LOG.md` (what was uploaded and what JLCPCB answered), `jlc-rotations.csv` and `jlc_final.py` (the rotation fixes applied to the CPL) |
| `release/revA/review/` | the review prints: 1:1 sheets, assembly drawings, copper layers, schematics, renders at A4 |
| `images/` | downscaled top renders for the README (left out of the engineering handover snapshots under `release/handover/`, as presentation, so the README's image links do not resolve inside a snapshot; they do in this repository) |

## State of the MESHSAT-830 generation

**Today (27 September 2026):** the foundations are incomplete and no board is ready for layout. The schematics of boards A, B, C, D, E and P carry the circuit corrections of 26 September 2026 and no committed layout carries them; the remaining blockers per board, and the step that closes each, are in `docs/CURRENT-EVIDENCE.md`. No routing campaign runs before its board's layout entry (`docs/EXECUTION-PLAN.md`). The rest of this section is the 7 September history.

The device set was ruled on 6 September 2026 (appendix 32.49 and 32.50), the fabric on 7 September (32.52: three slots, USB devices, k3s; not every device is a USB device, `docs/V2-SPEC.md` correction 6), and the five boards were generated from their generators the same day: A22 (the 14.4 V node, the charger, the rails, the outlet, eleven blind-mate sites, the D8 mezzanine site), B16 (three slots with their switches, hubs and drives, the Ethernet and HDMI switches, the radios), C7 (the backer ring with the RP2040 panel controller and the Pervasive Displays e-paper driver), D8 (the SA868 exciter, the amplifier leads, the USB audio path), E6 (the front end, the tracker, the pack entry, the sensor controller; the sensor board of the plan folded into it). The plan of that day was to route every board on a rented build host under `ecad/tools/routeflow.py` and to release a board when it was clean (0 unrouted, 0 hard DRC violations, the numeric gate passing), its deliverable folder landing in `release/revA/boards/`; `ecad/tools/check_contracts.py` then passed across the set (the 2x13 ribbons, the mezzanine harness, the EMCON chain, the four 5 V rails, the dock contacts). That reading is history: a board is now judged at the stage gates of `docs/EXECUTION-PLAN.md`, and no board has been released.

The JLCPCB cart of 3 September holds the previous generation and is not paid; its lines are rebuilt from the new deliverables when the owner declares the set final. On 25 September 2026 the owner ruled that the order folder `release/revA/order/` is to be rebuilt from the existing deliverable folders and quarantined, each order note carrying its board's readiness status, with nothing ordered and no cart line touched (decision 41, appendix 32.365). Parts fitted at the bench rather than by the assembler are listed per board in `ORDER-NOTES.txt` and in `docs/ASSEMBLY.md` section 9.

## Regenerating a board

The boards are generated by scripts, not drawn by hand. The pipeline runs headless on a rented build host (KiCad 9.0.9 with its Python bindings, Freerouting 1.9.0 built with a per-pass session, Java, Xvfb) driven by `ecad/tools/routeflow.py` with **one profile per board letter** in `ecad/tools/routeflow/<letter>.json`; everything that differs between boards is declared in `ecad/tools/boards/<letter>.json` (the phase, the pair classes and layers, the fanout nets, the finish stages) and the sequence lives once in `full.sh` and `finish.sh` (since 15 September 2026; before that there were 21 chain clones, 15 finish clones and 34 per-phase profiles).

1. `ecad/tools/full.sh <project dir> <letter>` writes the schematic (`gen_sch_<x>.py`, which also emits the netlist and the design-intent file), runs ERC, writes the outline and keep-outs (`gen_pcb_<x>.py`) and the placement, planes and locked rail copper (`gen_pcb_<x>3.py`), then the escapes of the fine-pitch parts, the pair pre-router (`pair_preroute.py`, every differential pair laid coupled before the router runs), the plane fanout, the same-net pin joins, the region-fit and placed-board DRC gates, and the placement predictor (`place_audit.py`); it stops with `PREROUTE-DONE OK` or `BLOCK`.
2. `python3 ecad/tools/routeflow.py run ecad/tools/routeflow/<letter>.json --phase <PHASE>` runs step 1, then Freerouting (single thread, the ground planes as power layers, a session written after every pass so a cut run keeps its best pass), judges the routed board and applies a bounded remedy per round; a run writes its provenance, its resolved configuration and a chained journal under `out/routeflow/<run>/`.
3. `ecad/tools/finish.sh` runs once per board: the knot repair, the dangling clean-up, the plane-pad vias, the pour stitching, the stub router for the last opens, the stitch and rail pruners, the return-current vias (a ground via beside every signal via), the quality pass, the pair length gate, the legend pass; every copper-editing pass runs under one guard (`guarded.sh`: snapshot, run, DRC, hard and unrouted against the board handed in, keep or restore). Then the routed-board gates: the fifteen-type hard DRC set, `check_pcb_<x>.py` with the return-path, decoupling and rail checks, `dc_drop.py`, `impedance_check.py`, `netlist_board.py`, `check_contracts.py`; then `finish_board.sh` cuts the deliverable folder and `verify_deliverable.py` reads it back.
4. `make_handoff.py` rebuilds `release/<rev>/order/` and `release/<rev>/review/` from the deliverable folders; `final_gate.py` re-reads every folder of the seven-board manifest with the contracts and the parts certification and fails closed on any of them.

The rules the tools hold are in `ecad/tools/tests/` (`python3 tools/tests/run.py` from `ecad/`; `tools/tests/run_code_only.sh` runs the same suite on a code-only archive). Prerequisites on the build host: KiCad 9.0.9 with `kicad-packages3d` (`kicad-cli` and `pcbnew` importable from `python3`), Java, the Freerouting 1.9.0 per-pass build (`tools/routeflow/cloud/onstart.sh` builds it from the v1.9.0 source; the stock jar is refused), Xvfb, `python3-numpy`, `python3-scipy`, and a venv with `build123d`, `ezdxf` and `matplotlib` for the CAD generators.

## Case

Peli 1450 without foam plus the 1450PF special application panel frame (CAD in `vendor/peli/1450/`). The frame window is 349.65 x 233.83 mm. By the session's case choices C1 and C6 (`docs/CASE-MARGINS.md` section 4), which the case generators carry since `c351115d`, the face plate is 377.2 x 263.0 x 3.0 on top of the frame over Peli's o-ring, on ten 6-32 screws into Peli's inserts, with the frame on four setting legs and the face top at 106.52 mm (the 7 September generation's plate was 365.5 x 249.5 x 3 on ten M3 at the frame's inserts, its top 101.4 mm above the cavity floor, the backer ring 10 mm under it); and the stack tops out at 49.5 mm at B16's top copper with the three coolers above it. The Xenarc monitor sits IN the plate with its glass level with the aluminium face, its body hanging into the void below (owner ruling 9 September 2026, appendix 32.85), the QMX HF unit rides in a printed tray on the lid's inner face (`release/case-2026-09-27/lid-tray-qmx-r2/`, sheets 14r2-1 to 14r2-3, which supersede the r1 tray and sheet 14 of that set: open across both end panels so every jack takes its plug, the unit lowered in from above and held by a screwed frame, on a lid plate bonded to the lid; its verification is open item %s), the pack lies in the east pocket under B16 (appendix 32.62; no pack is expected to fit the west pocket, `docs/V2-SPEC.md` correction 1), twelve arrestors at 59 mm on two RF entry plates are the antenna bulkheads (C2, C4; `ecad/tools/panel1450.py` is the single source of every face and wall position), and one connector plate between the hinge fairings outside the back wall carries the wall items (C3). The current case set, CAD, drawings and 1:1 templates, is `release/case-2026-09-27/`; `release/revA/case/` is the superseded 7 September set, kept as history and not to be made from; the interior numbers in design record 32.56 and 32.60.

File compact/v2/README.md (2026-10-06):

# MeshSat enclosure v0.6: LilyGO T-Beam Supreme + RockBLOCK 9704-SMA

**Status: cleared for PROTOTYPE printing. Not a final production release.**
See `AUDIT-RESPONSE.md` for how each audit finding (F01 to F15) was handled and what remains open.

Envelope (body + lid): **62.5 × 146.0 × 62.7 mm**; 154.0 mm long including the SOS guard.
With the MOLLE plate: 69.6 × 160.0 × 71.7 mm.

## Print in this order
| Step | File(s) | Material | Purpose / pass criterion |
|---|---|---|---|
| 1 | `coupons/meshsat-coupon_rails.stl` | PETG or ASA | The real 9704 PCB slides in with no flexing and no wobble. Otherwise change `rb_slot` (1.80) in the .scad. |
| 2 | `coupons/meshsat-coupon_rimlid.stl` | ASA | Inserts set flush; M3×8 screws close the lid onto the rim without bottoming; cord seats in the groove. |
| 3 | `coupons/meshsat-coupon_board.stl` + `print-stl/meshsat-separator.stl` + `print-stl/meshsat-lid.stl` | PLA ok | Real Supreme + 18650 seat on the separator. Lid closes without force. Buttons line up. OLED is centred in the window. |
| 4 | full set in `print-stl/` | PLA/PETG | Full prototype: assembly, wiring, dunk test |
| 5 | full set in `print-stl/` | **ASA** (orange) + TPU 95A | Only after steps 1 to 4 pass and the open items are closed |

| Part | Material | Orientation (already exported this way) | Notes |
|---|---|---|---|
| meshsat-body | ASA | open side up | 5 perimeters, ≥40 % infill; horizontal port holes may sag slightly, so deburr |
| meshsat-lid | ASA | outer face down | groove, pane pocket and hold-downs face up |
| meshsat-separator | ASA | flat underside down | 100 % infill |
| meshsat-membrane | TPU 95A | flange down, caps up | slow (20 to 30 mm/s) |
| meshsat-plungers ×3 | ASA/PETG | head down | |
| meshsat-retainer | ASA | flat | |
| meshsat-molle / -belt | ASA | body face down | tunnel roofs are 26.5 / 40 mm bridges: enable bridge settings or supports |

## Hardware
- **Lid:** 8× M3×8 socket head + 8× M3 heat-set inserts for a 4.0 mm hole, ≤ 5.7 mm long (pocket depth 7.0)
- **Carry plate:** 4× M3 heat-set inserts (same type) + 4× M3×8 countersunk
- **Button retainer:** 6× M2×6 self-tapping
- **9704 lock:** 2× M3×16 self-tapping, from above into the rail ends, after the board is slid in (fit before the separator)
- **Seal:** 2.0 mm silicone O-ring cord, ~450 mm. Groove 2.7 × 1.5 mm (77.6 % fill, 25 % squeeze). Join the ends with cyanoacrylate.
- **Foam:** 1.5 mm closed-cell foam: 1 strip ~15 × 70 under the 18650 holder, 4 pads 1.3 × 4 on the lid hold-downs (each compressed to 1.0 mm)
- **Window:** polycarbonate 24.0 × 38.0 × 2.0 mm (pocket 24.6 × 38.6 × 2.2), bonded with a neutral-cure silicone. Acetoxy (vinegar-smelling) silicone can craze polycarbonate.
- **Panel parts** (exact SKUs still open; check their cut-outs against the .scad):
  - 2× SMA female bulkhead pigtails with O-ring, Ø6.6 holes
  - IP67 panel USB-C, Ø16.2 hole; designed for a nut up to 20 mm across
  - M12 ePTFE vent, Ø12.3 hole on the right wall
  - 12 mm IP67 momentary switch, Ø12.2 hole, ≤ 20 mm deep behind the panel
- **Antennas:** Ground Control helical Iridium antenna (49 × 19 mm, SMA-M) + 868 MHz LoRa whip

## Assembly notes
1. RockBLOCK goes **component side down**. Slide it along the rails from the USB end until it hits the stop, then fit the two M3×16 lock screws.
2. Solder the harness wires directly to the 9704 header pins. There is ~3.9 mm under the pin tips, so Dupont housings won't fit. Anchor the bundle (adhesive tie mount in the free lower-bay area, y ≈ 25 to 55) so the solder joints carry no strain.
3. Fit the separator, then the foam strip, then the Supreme. Seat the PCB edges in the lips.
4. Fit the button membrane, plungers and retainer (6× M2×6) before closing.
5. Close the lid with even torque until it touches the rim. The rim is the hard stop, so don't overtighten.

## Electrical: open decisions (not designed here)
- **9704 power (F12):** Ground Control requires a battery supply to stay within 3.6 to 4.5 V on V_BATT. An 18650 drops below 3.6 V well before empty. Options:
  - (a) a 5 V boost converter feeding **V_IN+** (pin 15, 4.0 to 5.3 V, 500 mA); the lower bay has free space for one, y ≈ 22 to 56
  - (b) direct V_BATT with a firmware cutoff at about 3.7 V, accepting shorter runtime
  
  Use I_EN/I_BTD for start-up and shutdown. Connect all four 9704 grounds. Don't use the 9704's USB and header at the same time.
- **Co-location (F13):** Ground Control's installation page says the 9704-SMA Iridium certification assumes **no other transmitter in the same housing**, the qualified helical antenna with ≤ 0.5 dB feed loss, and the antenna ≥ 1 m above ground or metal. This design puts LoRa/BLE/WiFi in the same housing and adds a pigtail and bulkhead. **Get Ground Control's written position before a final build.**

## Rebuild and verify
`bash validation/build_and_check.sh` (OpenSCAD 2021.01+, Python: trimesh, numpy, scipy, manifold3d) regenerates every STL and reruns these checks:
- self-checks
- the clash check against the manufacturers' STEP meshes
- the mesh/printability report, including SHA-256 hashes

Results for this release are in `validation/build/`.

## Sources
- LilyGO T-Beam Supreme board STEP, DXF, schematic V3.1 and shell STLs: github.com/Xinyuan-LilyGO/LilyGo-LoRa-Series, commit 5e2da3f. © LilyGO; included for reference only.
- RockBLOCK 9704-SMA (2A) STEP, mount STEP + drawing, Maxtena antenna STEP: docs.groundcontrol.com/iot/rockblock-9704/hardware. © Ground Control; included for reference only.
- `reference-cad/meshes/*.stl` are tessellations of those STEP files, used for the assembly view and the clash check.

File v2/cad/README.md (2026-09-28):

# v2/cad: the case set's editable sources and how to regenerate them

MESHSAT-1357, 27 September 2026. Prototype design: nothing in this folder has been made, bought or fitted. The released copies are
`v2/release/case-2026-09-27/`; the files here are the authority, the release folder is an immutable copy of what they produced.

## What is here, and what is current

| File | What it is | Current? |
|---|---|---|
| `../ecad/tools/panel1450.py` | **The single geometry source** of the case set: Peli's figures the arrangement derives from, the face plate (C1), the setting legs (C6), the stack, the connector plate and its six items (C3), the RF entry plates and the twelve arrestor sites (C2, C4), the QMX tray's place (C5), the pack block's place. Plain Python; board C's gate, the face budget and every file below read it. | current |
| `zstack.py` | Reads the committed KiCad boards (the file each board's routeflow profile names, and board E5) with the standard library: outlines, holes, thickness, and every footprint's side, plan rectangle and height (its own library model's, from `zstack-models.json`, or a declared class). A library model is a nominal body, so where a worst-case chain takes a part's height the maker's maximum is read off its sheet and carried beside it (`MAKER_MAX`: U51, STM32H753VITx in LQFP-100, 1.60 by ST's DS12117 Rev 9 Table 217, whose typical 1.50 is the model's). Writes `zstack.json`; prints the Z stack and the bays. | current |
| `zstack.json` | The board reading: each board file with its sha256, its parts with heights and their sources (and `height_max` where `MAKER_MAX` gives one), the bays, and `b16_envelopes`, which `panel1450.B16_TALL` loads for the face gates on first use. **Required, never replaced:** without it `panel1450.B16_TALL` raises `ZstackMissing`, so board C's gate reads INCONCLUSIVE instead of passing on a weaker list; a tree a gate runs in must carry it (`drafts/hc7/stage_chain.sh.patch` stages it into chain trees). | current (regenerate when a board changes: the test says so) |
| `zstack-models.json` | The KiCad 9 library models the boards name (kicad-packages3D tag 9.0.9): sha256 and bounding box of each, SUBSTITUTE where the named file is missing from the library, the error where neither exists. | current |
| `model_bbox.py` | Writes `zstack-models.json` (needs the network and the CAD set below). | current |
| `face_plate.py`, `plate_drawing.py` | The face plate (C1): STEP, STL, DXF (layers OUTLINE, THROUGH, POCKET_1MM, REBATE_2MM_TOP, RELIEF_0.8MM_UNDERSIDE, STANDOFF_M3), marking SVG; its dimensioned drawing (sheet 1). | current |
| `frame_leg.py` | The four setting legs (C6), their printed locator and the centring wedges: STEP, STL, the leg's DXF profile. | current |
| `connector_plate.py` | The back wall's connector plate (C3) and its gasket: STEP, STL, DXF (seen from outside). | current |
| `rf_entry_plate.py` | The two end walls' RF entry plates (C4) and their gaskets: STEP, STL, DXF per wall (seen from outside). | current |
| `case_drawings.py`, `drawing_kit.py` | Sheets 2 to 14: frame and legs, connector plate, RF entry plates, the Z stack, the case in plan, the seven board envelopes, and the QMX lid tray with its place on the lid (sheet 14, added 27 September 2026 by the layer 7 fixer c7). Every sheet names its inputs by sha256 and labels the margin rows its features enter (MET or OPEN, read from `../vendor/peli/1450/frame_seat.out`). | current |
| `../ecad/tools/case_wall_cutouts.py` | The 1:1 marking templates (back wall, east wall, west wall) and check prints (connector plate, both entry plates, the face plate on A3). | current |
| `case_geometry_check.py` | The drift checks `../ecad/tools/tests/test_case_geometry.py` runs: board identity, the face gates' coverage of board B, the face basis against `frame_seat.out`, `frame_seat.py` against its record, the makers' maxima on board parts, the worst-case reads of `frame_seat.py` (a worst-case chain takes `height_max`, never a model's nominal height), a release folder against its manifest. | current |
| `build_case_release.sh` | Regenerates the whole case set into a folder, copies the margins it is labelled with and writes its manifest. | current |
| `case_manifest.py` | Writes a release folder's `MANIFEST.sha256` (stdlib); run it again after the folder's README.md is written. | current |
| `lid_bracket_qmx.py` | **Superseded by the r2 tray below.** The QMX lid tray (C5) of r1: STEP and STL of the part of 9 September 2026, unchanged; its numbers are module constants and its place across the case (`PLACE_Y`, Y -51.5 to 71.5) sits beside them, so sheet 14 reads the part and `panel1450.QMX_TRAY_X` (X 102.0 to 171.0) instead of retyping them. Importing it builds nothing. **Its fit to the unit is OPEN** (the QMX's jacks are on both end panels and the tray is notched at one end only; `v2/docs/CASE-FIT-UNCERTAINTIES.md` section 3). | superseded (27 Sep 2026) by `lid_tray_qmx_r2.py`; kept because the released r1 files and sheet 14 were made from it |
| `lid_tray_qmx_r2.py` | The QMX lid tray r2 (S-63, EQ-24; second pass of 27 to 28 Sep 2026): the tray, its retaining frame and its aluminium lid plate from the maker's dimensions (`../vendor/qrp-labs/`), open at both end panels, the unit lowered in from above and held under the screwed frame, top face out with its right panel toward the hinge; STEP, STL, the plate's DXF. `elements()` is the one table of solids the parts are built from and the check and the sheets read. Its jack, knob and LCD places are the scaled figures of `../vendor/qrp-labs/qmx-figures.out` (`measure_qmx_figures.py`); its east edge stays at `panel1450.QMX_TRAY_X[1]` (C5, M19 unchanged) and its place (`PLACE_X`, `PLACE_Y`, `SPAN_X`, `SPAN_Y`) sits beside the part. Importing it builds nothing. | current |
| `lid_tray_qmx_r2_check.py`, `lid_tray_qmx_r2_drawing.py`, `build_lid_tray_r2.sh` | The r2 record: each jack's admitted plug body and the leads' room (A); the face room, every row from the deepest solid over each face part, with the part's height from its maker's sheet and the set's own allowances (B); the pads (C); the load case and every retention link (D); the fitting, the unit at its largest and the frame swept along their way in against every solid (E), with two controls that must fail (the first pass's tray and way in, the first pass's face-room row). With `--solids`: the table against the built solids, the unit, the plug bodies and the knobs in place, and both ways in position by position. Sheets 14r2-1 to 14r2-3, and the script that builds all of it into `lid-tray-qmx-r2/`. `../ecad/tools/tests/test_lid_tray_qmx_r2.py` checks the numbers and both controls without the CAD set. | current |
| `pack_4s.py` | The rigid 4S pack box of 7 September 2026. **Superseded**: it fits no pocket (adjudication A06, W4-F3); the ruled pack is a shrink-wrapped 4S3P block (D-06) whose hold-down is not designed (S-27, CON-006). Kept for the record only. | superseded |
| `battery_module.py` | The retired twelve-cell module. | superseded |
| `float_clamp.py` | The dock's float nest for the SMP-MAX plugs: its 16 mm nests overlap at the 14 mm site pitch; one clamp bar (R4E-07) is owed. | not current |
| `render/` | The concept render scene of 5 to 9 September 2026 (Blender 4.2 on a GPU host). It draws the superseded face (rim 109.4, plate under the ring), the Amphenol couplers at Z 88 and the old connector plate; its images are illustrations of that state, not of this set. Not regenerated here. | superseded for measurement |
| `stack-heightmap.json` | The height map of 5 September 2026 (from the render scene). Superseded by `zstack.json`. | superseded |

## Regenerate

Host: any Linux x86_64 (the release was made on Ubuntu 24.04.5 LTS with Python 3.12.3). No KiCad, no Blender, no GPU and no particular
host is needed; only `model_bbox.py` needs the network.

```
python3 -m venv .venv-cad
.venv-cad/bin/pip install -r v2/cad/requirements-cad.lock      # the exact set; requirements-cad.txt names the six top-level pins
v2/cad/build_case_release.sh /tmp/case-out                      # PY=.venv-cad/bin/python by default
REFETCH_MODELS=1 v2/cad/build_case_release.sh /tmp/case-out     # also re-fetch the KiCad library models (network)
```

The standard-library parts run on any Python 3.8 or later without the venv:

```
python3 v2/cad/zstack.py --report                 # the Z stack and the bays, from the committed boards
python3 v2/ecad/tools/z_budget.py                 # the face budget (M1), from panel1450.py
python3 v2/vendor/peli/frame_seat.py              # every case margin (70 rows) and its verdict
python3 v2/cad/case_geometry_check.py             # the drift checks
python3 v2/ecad/tools/tests/run.py case_geometry  # the same, with the defective fixtures
python3 v2/cad/lid_tray_qmx_r2_check.py           # the QMX lid tray r2's record (add --solids in the venv for the checks on the solids)
python3 v2/ecad/tools/tests/run.py lid_tray_qmx_r2
```

The QMX lid tray r2 alone, into `<out>/lid-tray-qmx-r2/` (with the venv): `PY=.venv-cad/bin/python v2/cad/build_lid_tray_r2.sh <out>`;
read the three page images it leaves in `<out>/.lid-tray-qmx-r2-readback/` before a release takes the folder, write the folder's
`README.md`, then `python3 v2/cad/case_manifest.py <out>/lid-tray-qmx-r2 --base <commit>` for the set's own `MANIFEST.sha256`. The r2 set is a folder
beside the case release's files, with its own manifest: the release's `README.md` and `MANIFEST.sha256` are not edited for it.

STEP and PDF files carry time stamps: two builds of the same sources differ in those bytes. Compare geometry (the printed sizes and
volumes, the DXF entities) and the drawings, not the file hashes; the release's `MANIFEST.sha256` identifies the files as released.

## How a change flows

1. Change a number in `panel1450.py` (or a board file, then run `zstack.py --json v2/cad/zstack.json`).
2. Run `frame_seat.py`; if a figure or verdict moves, update `v2/docs/CASE-MARGINS.md` and commit the new `frame_seat.out` with it.
   `frame_seat.py` reads its design numbers from `panel1450.py` and its board inputs from `zstack.json` from the change that follows this
   release (the frame_seat.py draft of MESHSAT-1357, 27 September 2026); until that lands it types them, and `case_geometry_check.py`'s
   `literal_inputs` and `worst_case_reads` name the two typed inputs (U51's height, typed as 1.6 from the LQFP class, which is ST's
   maximum 1.60 the draft reads from `zstack.json`; and a six-part hand list of B16's tall parts, which misses the E72 module U14).
3. Run the drift checks, then `build_case_release.sh` into a NEW release folder `v2/release/case-<date>/`, write its README.md (source
   revision, inputs by sha256, what it supersedes, what is open), run `python3 v2/cad/case_manifest.py v2/release/case-<date>/` last, and
   mark the previous folder superseded in its README. A release folder is never edited in place.

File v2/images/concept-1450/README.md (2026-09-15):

# Concept renders, the kit in the Peli 1450 (rendered 7 September 2026, eighth set: the MESHSAT-830 board set)

> **15 September 2026, set nine (`set-nine/`, 18 views):** the monitor in set eight below stands 28.7 mm proud of the face plate,
> a scene defect corrected on 9 September (design record 32.85: the Xenarc sits IN the plate with its glass level with the
> plate's top face, held to 1 mm at most). Set nine renders the corrected scene with the boards as they stand on 15 September
> (A32, B19 placed, C17, D11, E9, E5, P4); read `set-nine/README.md` for its views. The images below are set eight and are
> superseded where they show the face.

Concept illustrations of the V2 kit as designed on 7 September 2026 (design record 32.49 to 32.61): the Peli 1450 with the 1450PF frame, the 3 mm aluminium face plate with the Xenarc 709GNK monitor lying on it, the backer ring C7 under it, the RA30H1317M1 amplifier module on the plate's underside, the rod stack of A22 (with the D8 mezzanine) and B16 (three Compute Module 5 slots with their coolers, the M.2 cards and drives, the LimeSDR bay, the RockBLOCK, the radios), the dock strip E6 with the raised block E5 and the eleven blind-mate float clamps, the eleven SMA couplers at Z 88 in the end walls, the connector plate on the back wall and the QMX HF unit in its tray on the lid. The BB-2590/U is not drawn: its place is the open ruling of 32.60 item 7 and 32.61 item 7. Blender 4.2 Cycles on an H100 box, the boards from the released KiCad projects (`kicad-cli pcb export glb` with the library models), the case from Peli's drawing 1451-931, the makers' STEP files for the modules, stand-in shapes for the rest. Nothing has been built; every picture is design intent.

Every image carries rulers (white bars, 10 mm ticks, numerals every 50 mm) along the case's edges on the ground and standing at the front corners, a 50 mm floor grid, and a title strip with the view name.

## The inside

**stack-no-face-top**: the stack from above with the face plate and backer removed: B16 with the three Compute Modules and their coolers, the NVMe drives and the cards, the LimeSDR in its bay, the RockBLOCK, the LG290P, the E22 and the two E72, the panel ribbon and the HDMI cable.

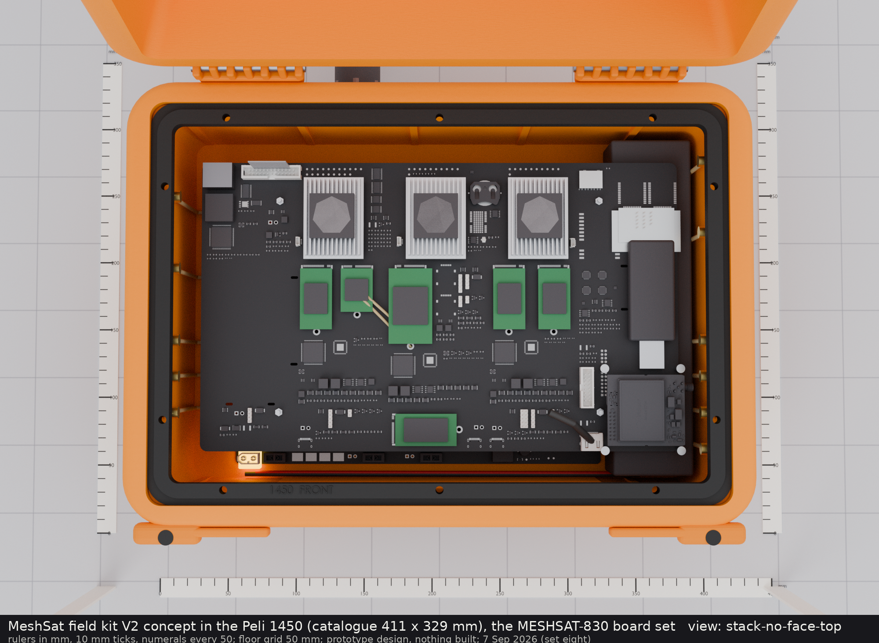
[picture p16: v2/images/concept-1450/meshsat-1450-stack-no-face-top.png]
stack-no-face-top


**stack-no-face**: the stack without the face, three-quarter view.

stack-no-face

**stack-no-face-east**: the same from the east end.

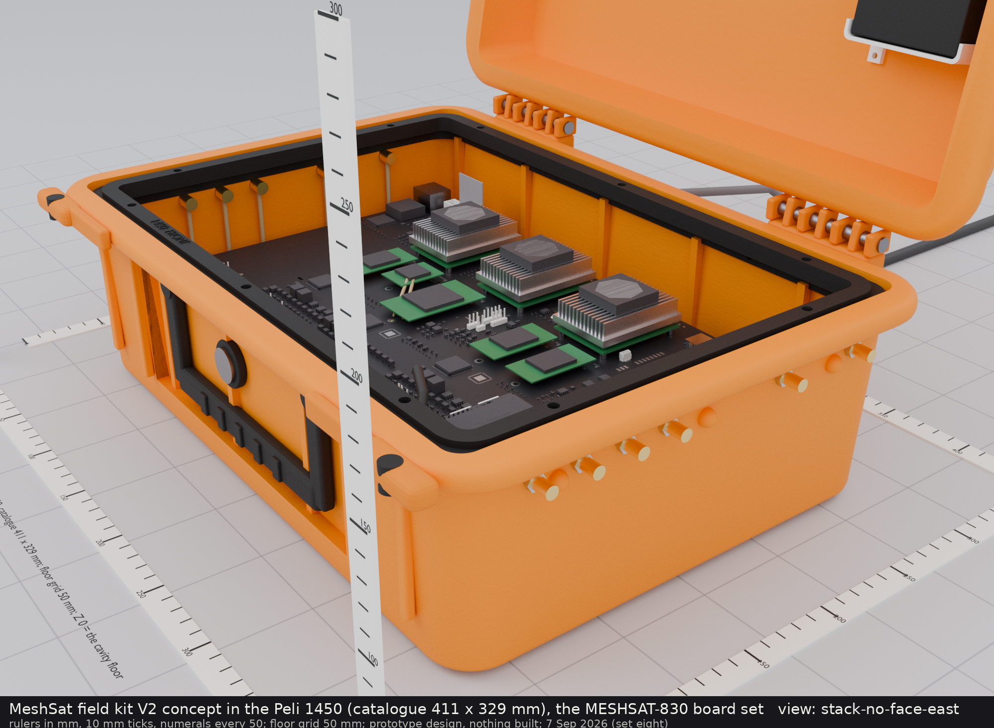
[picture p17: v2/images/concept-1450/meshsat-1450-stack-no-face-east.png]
stack-no-face-east


**stack-no-face-back**: the same from the hinge side.

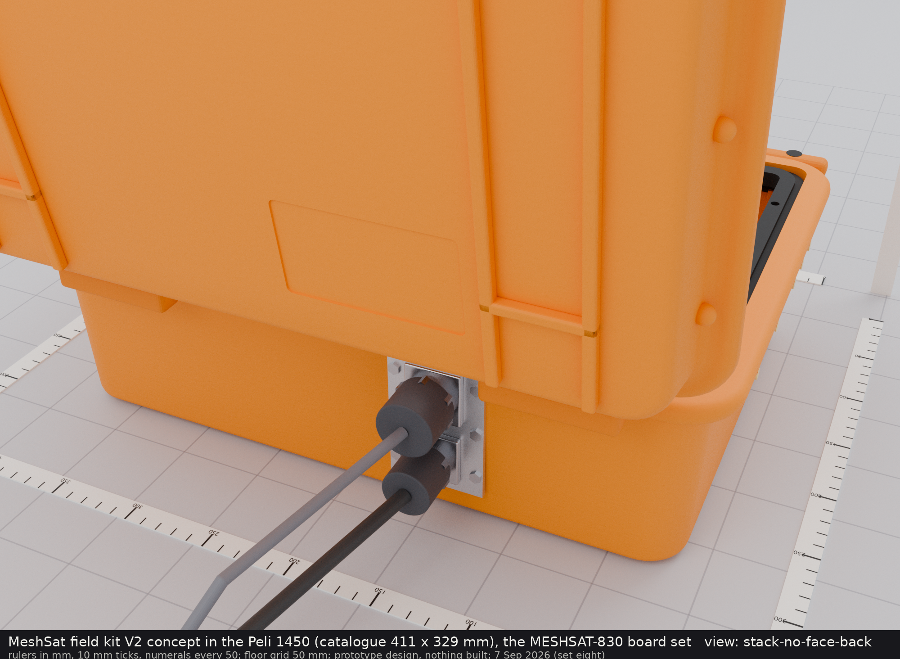
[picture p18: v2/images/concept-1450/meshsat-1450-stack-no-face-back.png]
stack-no-face-back


**level-b16**: B16 on top of the stack.

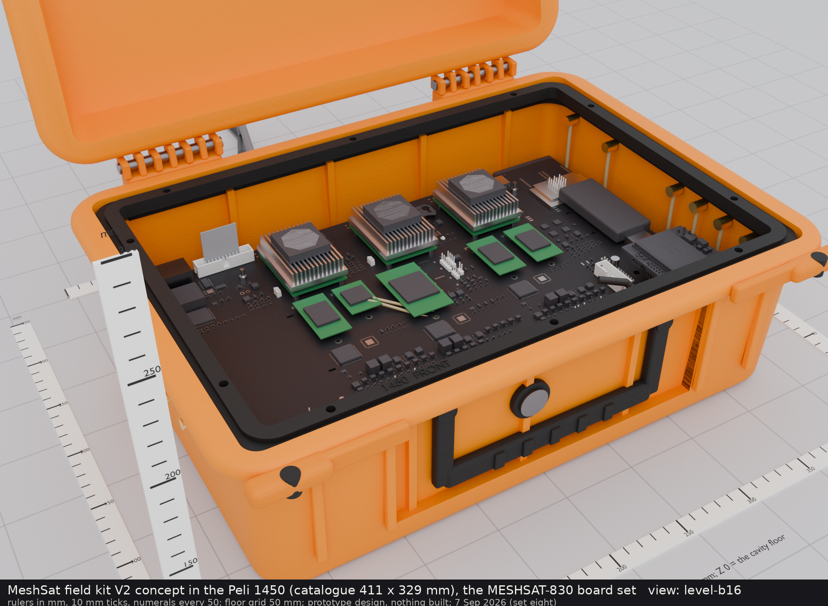
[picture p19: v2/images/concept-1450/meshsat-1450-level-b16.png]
level-b16


**level-d8**: B16 lifted away: D8 on its standoffs on A22, the SA868, the relay and filter, the leads to the amplifier.

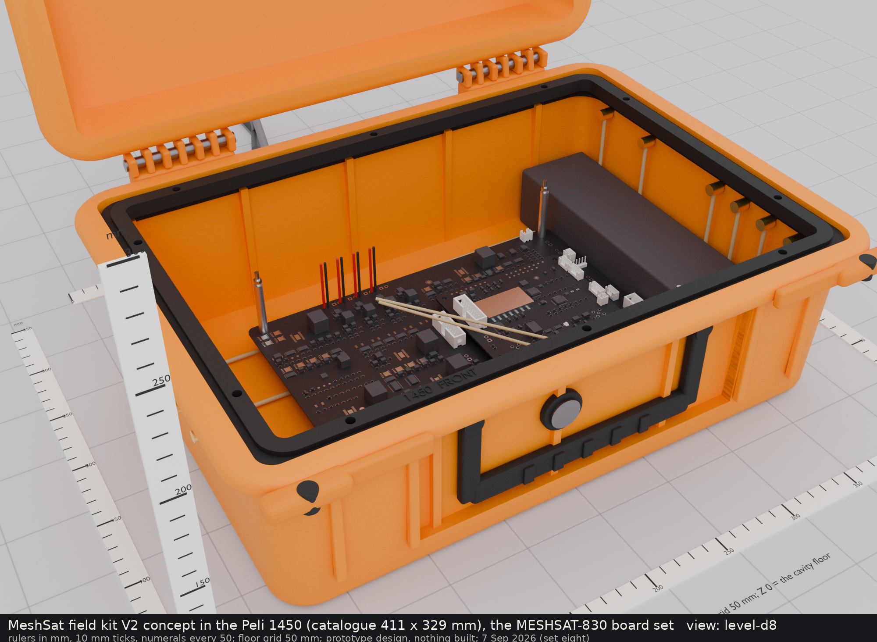
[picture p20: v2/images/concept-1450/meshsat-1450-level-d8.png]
level-d8


**level-a22** and **level-a22-top**: A22 alone on the rods: the converters, the charger, the eleven SMA jacks over their blind-mate receptacles, the dock contacts.

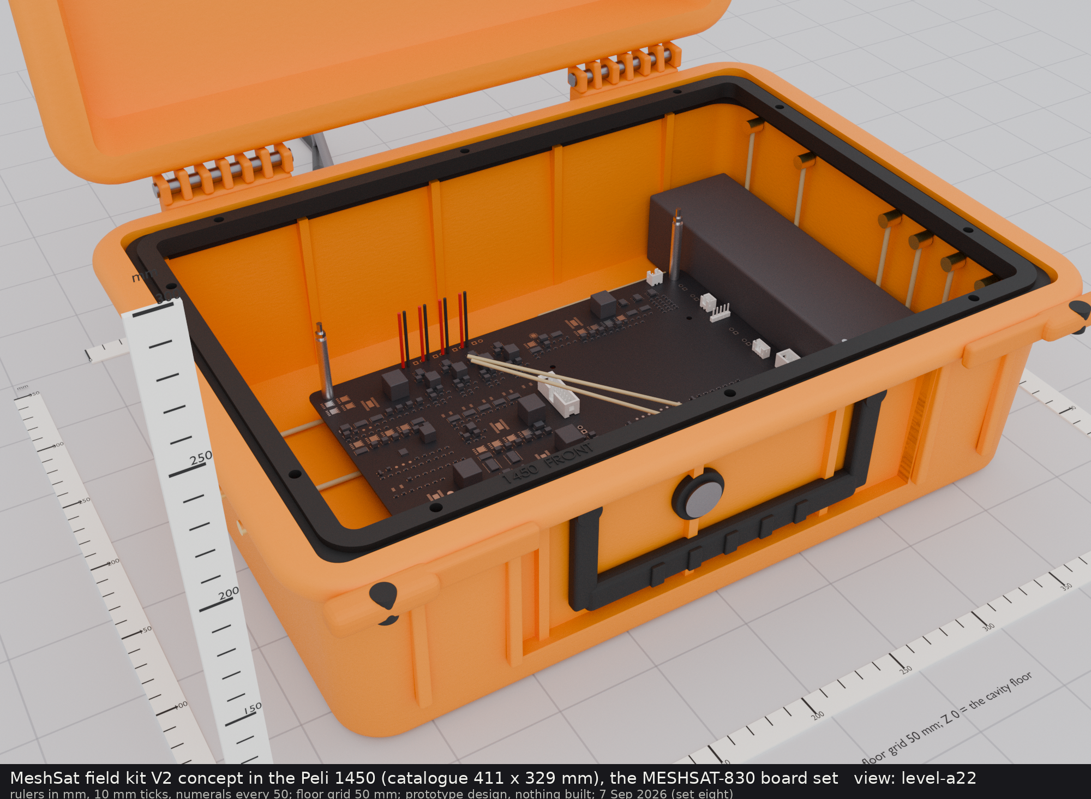
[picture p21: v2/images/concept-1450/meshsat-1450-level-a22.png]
level-a22


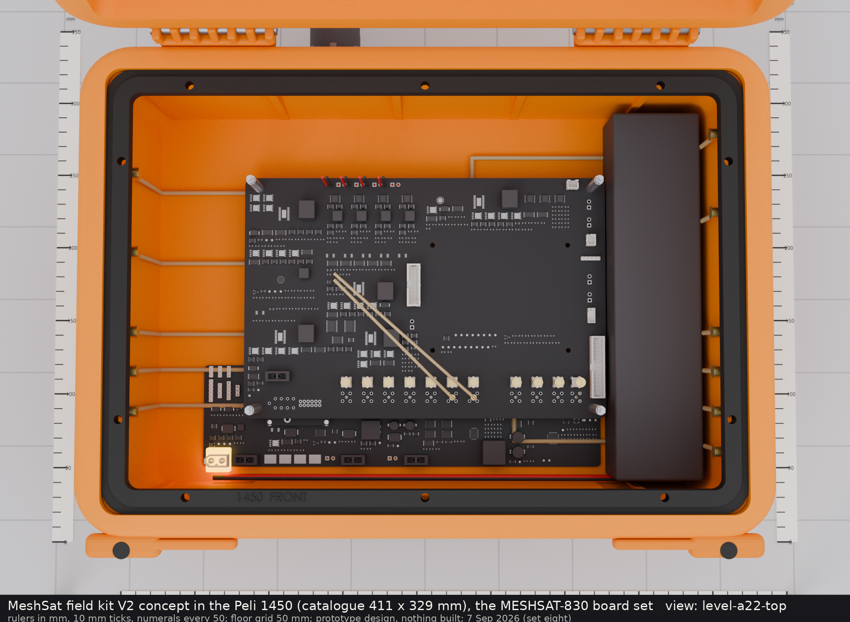
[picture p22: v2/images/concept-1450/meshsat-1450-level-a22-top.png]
level-a22-top


**level-dock** and **level-dock-top**: the empty case floor: the dock strip E6 with the block E5, the eleven float clamps and their pigtails to the end walls, the sensor headers.

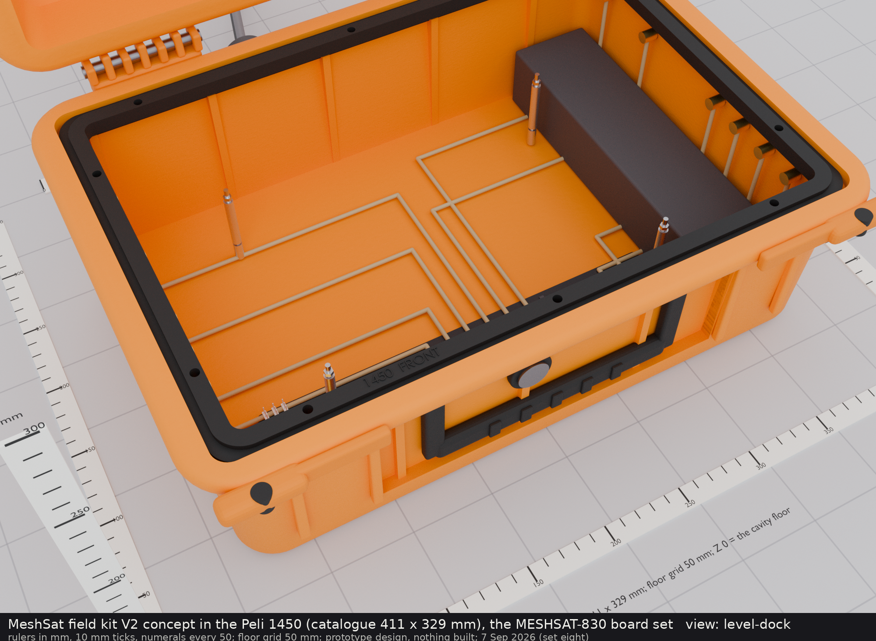
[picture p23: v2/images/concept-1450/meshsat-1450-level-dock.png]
level-dock


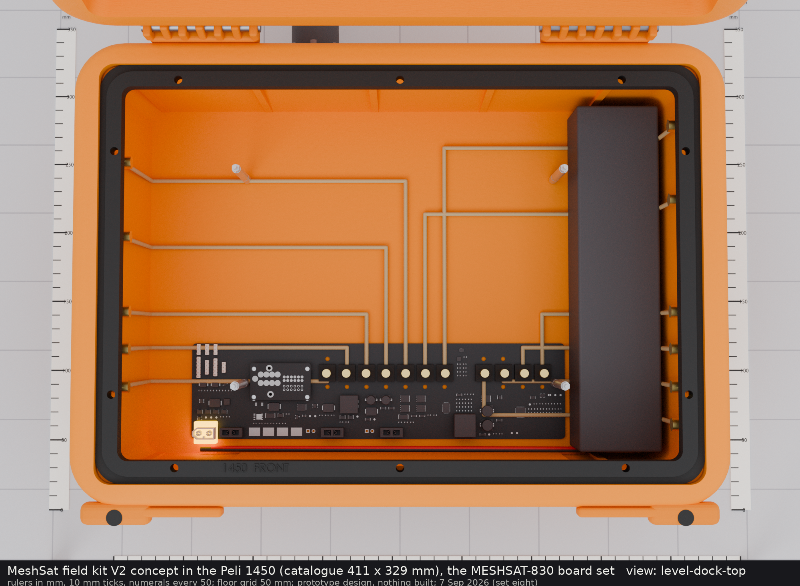
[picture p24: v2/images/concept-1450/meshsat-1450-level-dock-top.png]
level-dock-top


**dock-joint** and **dock-joint-a22**: the front wall removed: the float clamps and the right-angle plugs on the dock strip, then A22 mated on them.

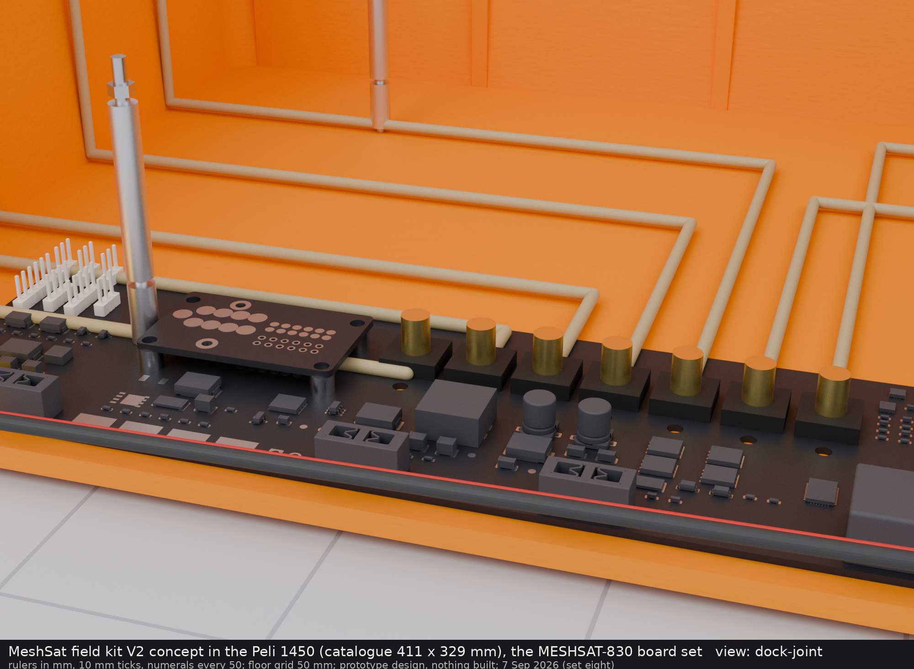
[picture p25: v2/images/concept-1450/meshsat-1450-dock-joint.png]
dock-joint


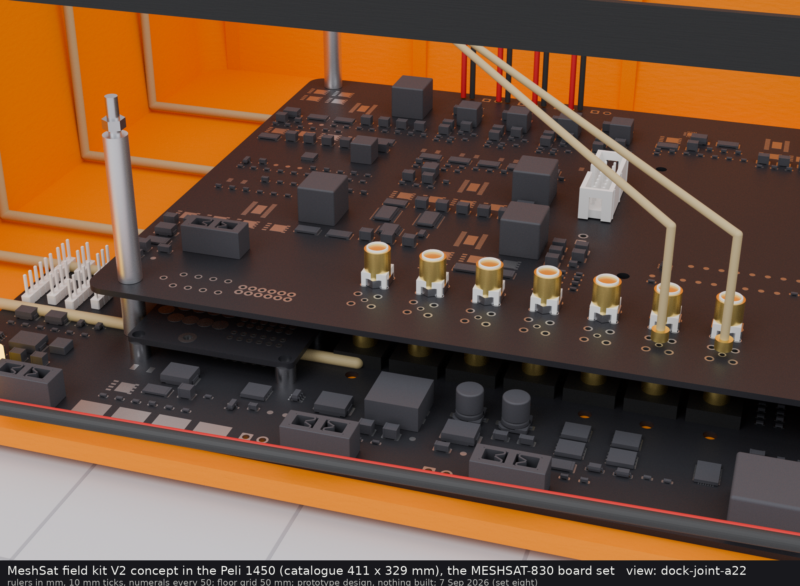
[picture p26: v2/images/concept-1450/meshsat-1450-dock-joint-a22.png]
dock-joint-a22


**cutaway** and **cutaway-east**: the front wall cut away and the face lifted on its ribbon: the whole stack in place.

cutaway

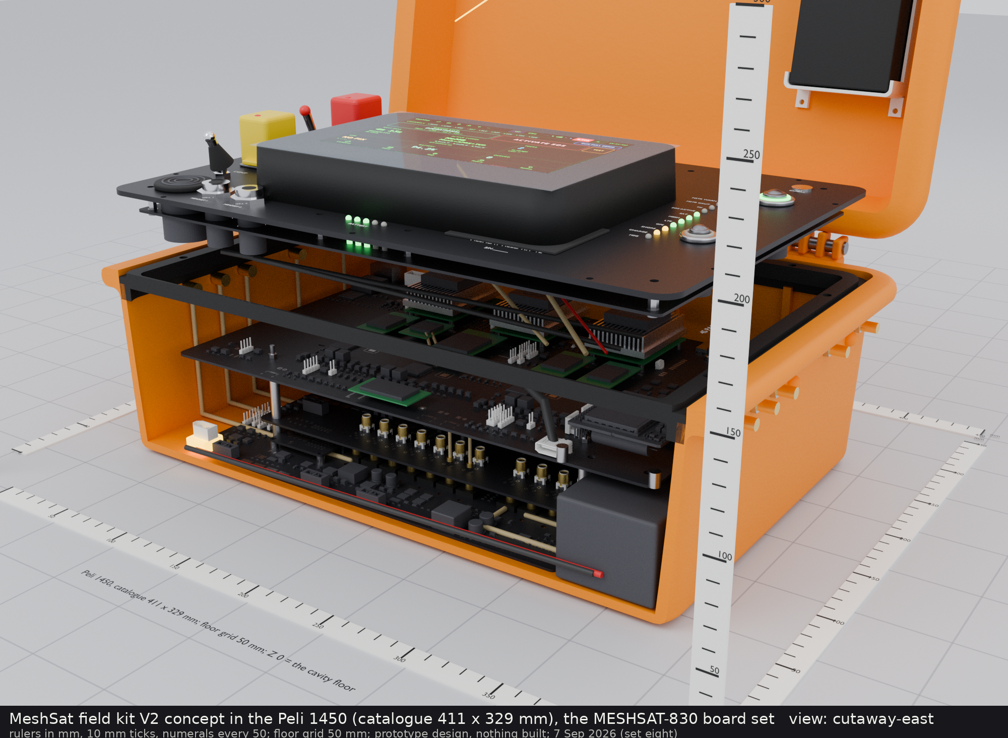
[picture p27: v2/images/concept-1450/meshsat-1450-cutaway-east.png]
cutaway-east


**west-wall-inside** and **east-wall-inside**: the end walls from inside: the five and six couplers at Z 88 with their pigtails down to the dock clamps.

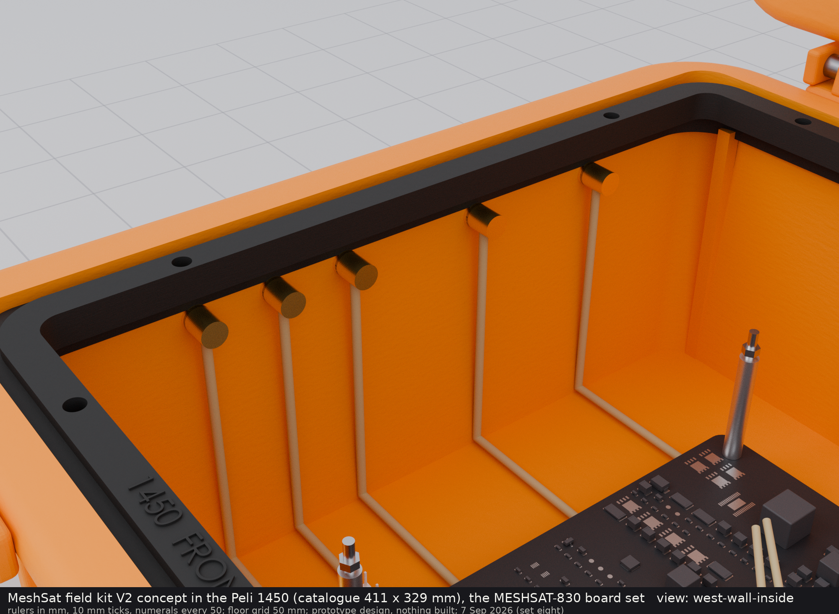
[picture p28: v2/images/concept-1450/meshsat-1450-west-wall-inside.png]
west-wall-inside


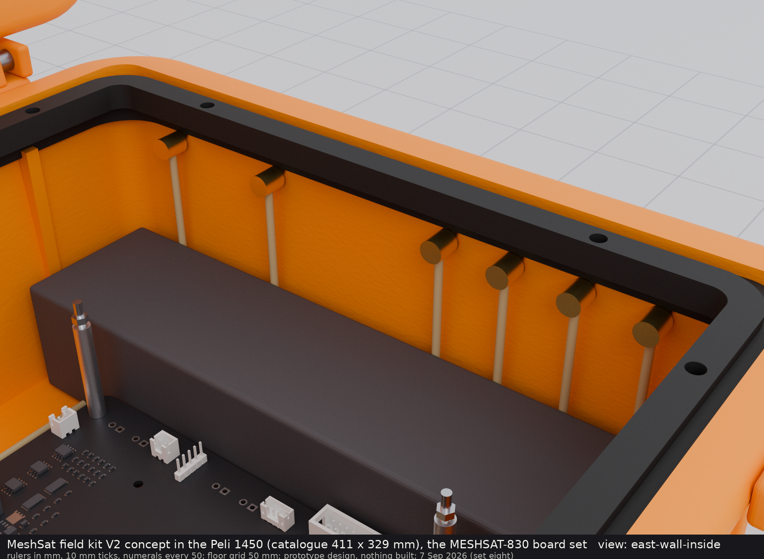
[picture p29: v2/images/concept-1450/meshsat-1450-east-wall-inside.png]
east-wall-inside


## The face

**top-face**: the face from above: the Xenarc monitor with the kiosk page, the e-paper with the QR code, the switch column, the indicator column, the headset jacks, the camera and light sensor windows, the legends.

top-face

**face-detail-left** and **face-detail-right**: the two switch corners.

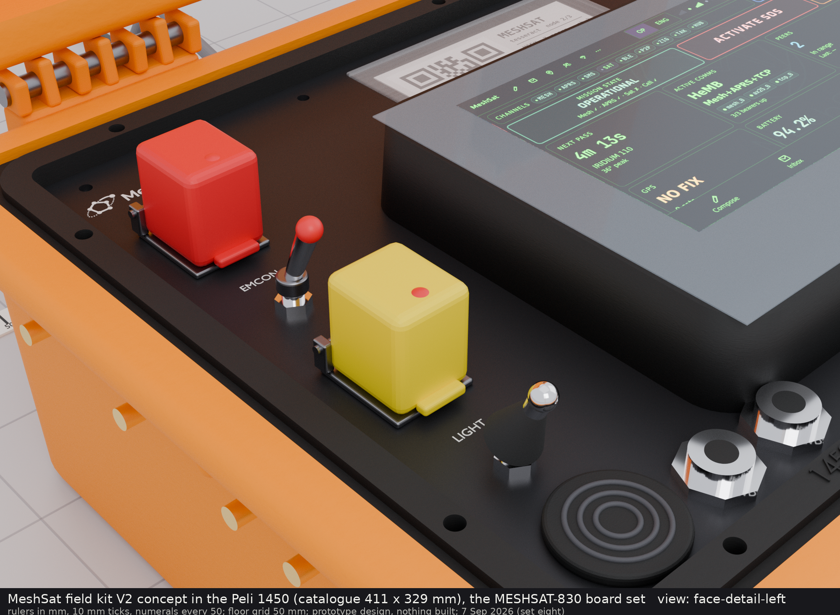
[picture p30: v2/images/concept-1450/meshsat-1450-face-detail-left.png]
face-detail-left


face-detail-right

**face-underside** and **face-underside-top**: the plate lifted 150 mm on its ribbon: the backer ring C7 on its eight standoffs, the monitor's connector block through the plate, the e-paper flex, the LEDs under the light guides.

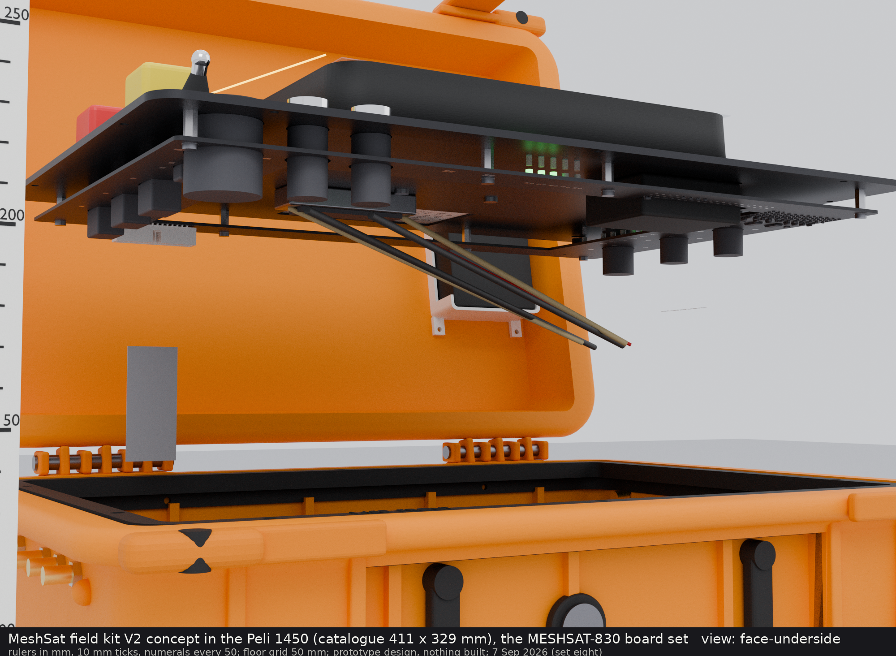
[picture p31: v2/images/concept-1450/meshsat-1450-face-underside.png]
face-underside


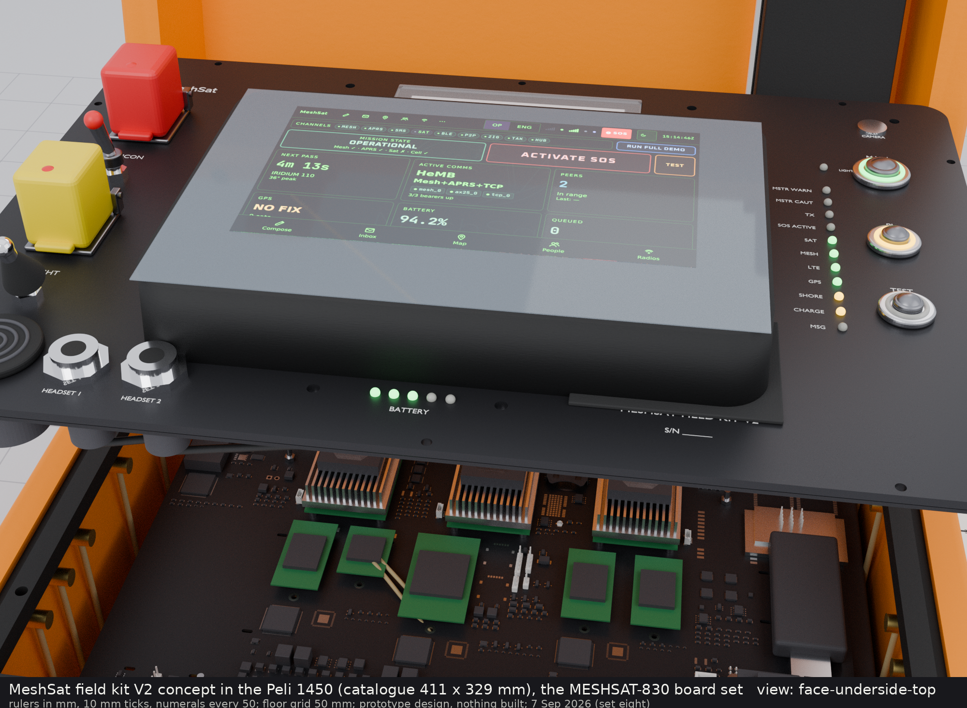
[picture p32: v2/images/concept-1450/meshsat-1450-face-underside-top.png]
face-underside-top


**face-pa-underside**: the amplifier module bolted flat under the plate on its two nuts, its leads down to D8.

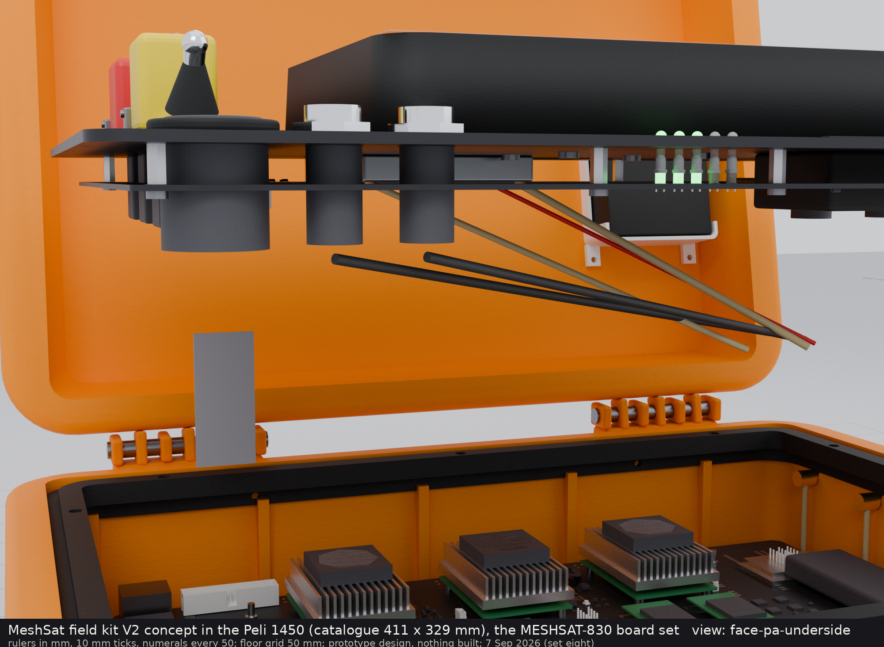
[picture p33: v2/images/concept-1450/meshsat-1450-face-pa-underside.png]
face-pa-underside


**lid-inside**: the open lid's inner face: the QMX tray over the right strip with the unit strapped in.

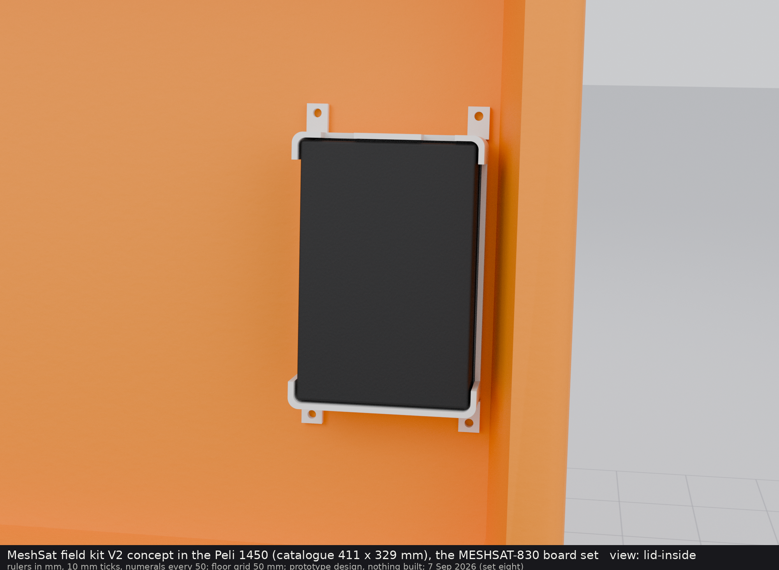
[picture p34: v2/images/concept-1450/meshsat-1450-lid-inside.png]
lid-inside


## The case

**az000-el40-open** to **az315-el40-open**: eight orbit views with the lid open, elevation 40 degrees.

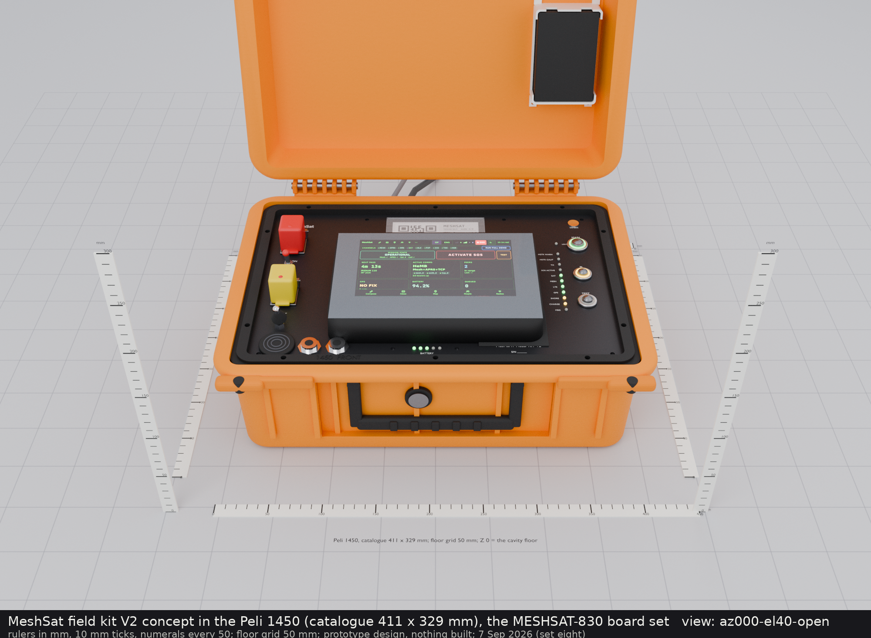
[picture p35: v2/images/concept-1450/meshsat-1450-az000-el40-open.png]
az000-el40-open


az045-el40-open

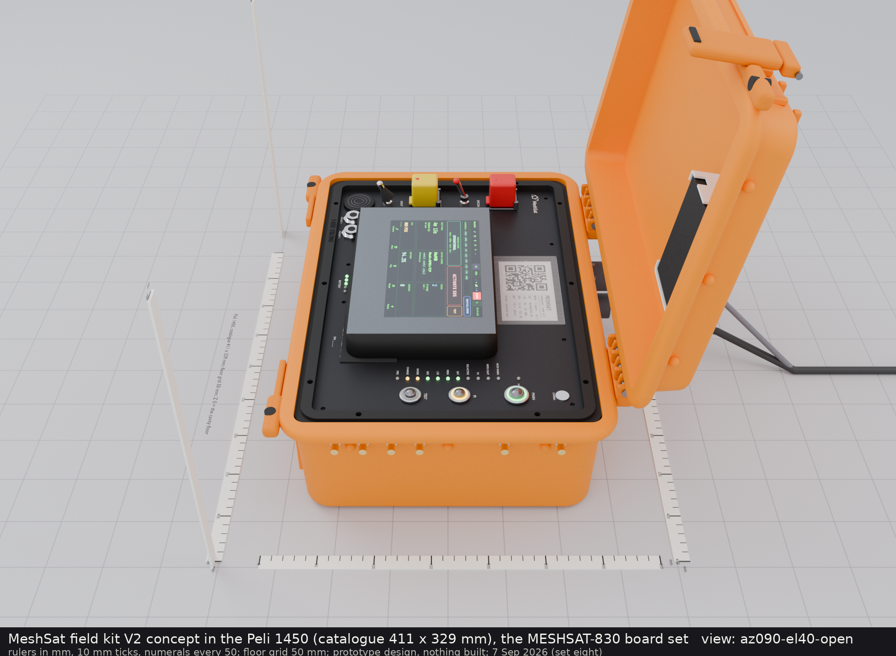
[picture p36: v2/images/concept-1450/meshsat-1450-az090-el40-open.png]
az090-el40-open


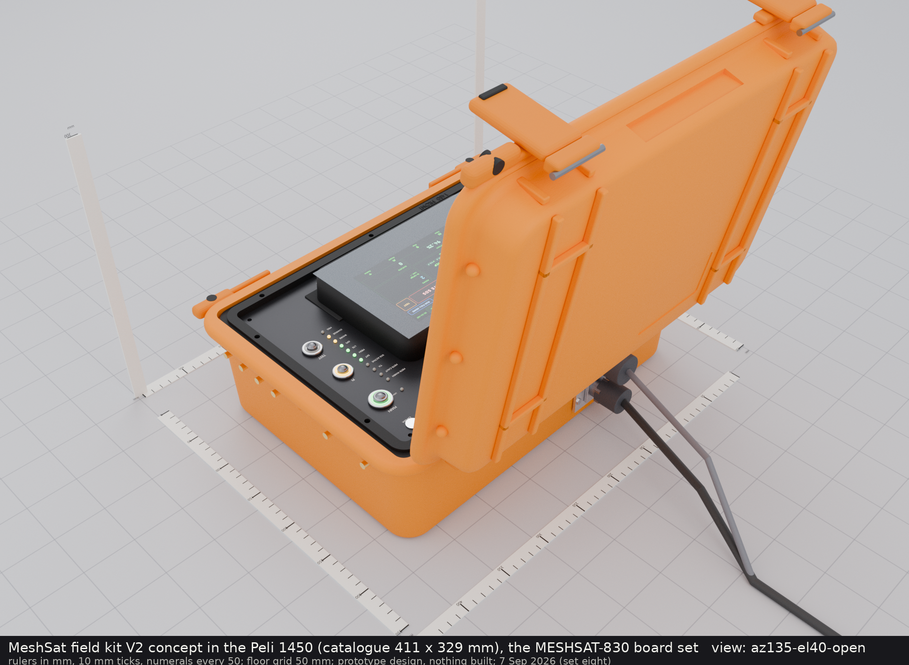
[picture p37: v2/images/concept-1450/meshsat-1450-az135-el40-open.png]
az135-el40-open


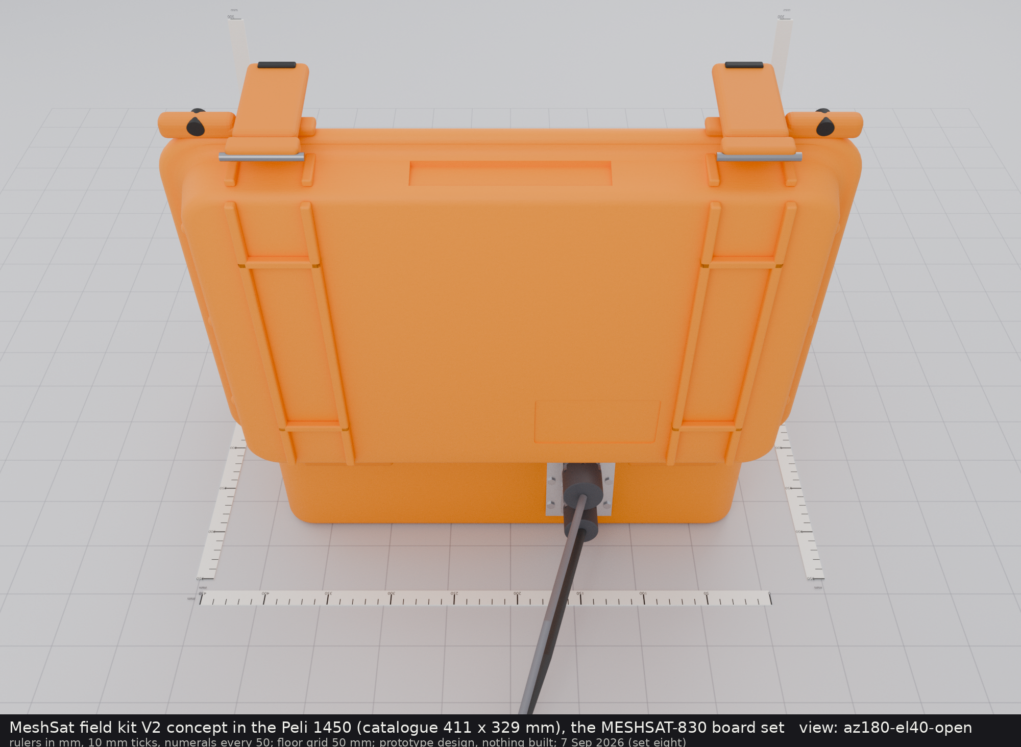
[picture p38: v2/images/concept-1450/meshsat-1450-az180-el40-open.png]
az180-el40-open


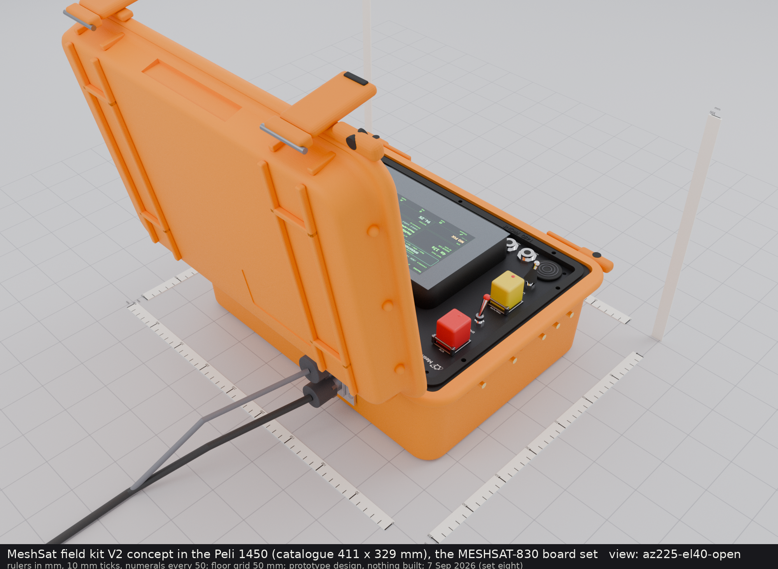
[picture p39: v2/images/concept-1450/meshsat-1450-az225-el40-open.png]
az225-el40-open


az270-el40-open

az315-el40-open

**az135-el40-open-nocables**: the same view without the external cables.

az135-el40-open-nocables

**az000-el20-closed** to **az270-el20-closed**: four views closed for transport, elevation 20 degrees.

az000-el20-closed

az090-el20-closed

az180-el20-closed

az270-el20-closed

**west-wall**, **east-wall**: the end walls from outside with their coupler rows and legends.

west-wall

east-wall

**back-wall**, **back-wall-nocables**, **connector-plate**: the back wall with the connector plate, both cables plugged and unplugged.

back-wall

back-wall-nocables

connector-plate

**antennas-az045**, **antennas-az315**, **antennas-az225**, **antennas-top**: the kit with every antenna fitted (the VHF whip, the HF wire kit's feed, the WiFi and P2P whips, the GNSS puck on the ground beyond the west wall, the SDR whip, the 5G stubs, the Iridium helical, the LoRa whip).

antennas-az045

antennas-az315

antennas-az225

antennas-top

## Disassembly in five pictures

**assembly-1-closed**, **assembly-2-lid-open**, **assembly-3-plate-off**, **assembly-4-stack-out**, **assembly-5-dock**: the sequence of `docs/ASSEMBLY.md`: closed; lid open; the face plate assembly lifted and set down east; the rod stack lifted off the blind-mate joint and set down west; the empty case with the dock.

assembly-1-closed

assembly-2-lid-open

assembly-3-plate-off

assembly-4-stack-out

assembly-5-dock

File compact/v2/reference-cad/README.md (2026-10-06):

# Reference CAD for the compact v2 enclosure

Third-party models and drawings the enclosure was registered against, kept so the design can be checked against the same files later. **They are not covered by this repository's licence.** Each file belongs to its maker under that maker's terms and is kept here as reference material for the design record. If you hold the rights to one of these files and want it removed, open an issue and it goes.

| Folder | Source | Used for |
|---|---|---|
| `lilygo-t-beam-supreme/` | LILYGO T-Beam Supreme: the board STEP (`T-Beam-Supreme-board.stp`), the V3.0 DXF, the V3.1 schematic PDF, and under `lilygo-shell/` the three STL files of LilyGO's own shell; from github.com/Xinyuan-LilyGO/LilyGo-LoRa-Series at commit 5e2da3f. © LILYGO | the board's registration in the upper bay (PCB 1.0 mm, the tallest top-side part, the three side buttons' actuator faces, the OLED window), and the 18650 holder envelope, which the STEP does not carry and the shell does |
| `groundcontrol-rockblock-9704/` | Ground Control RockBLOCK 9704-SMA: the mount STEP (Rev A) and the Maxtena helical antenna STEP (100-00003-02 Rev B); from docs.groundcontrol.com/iot/rockblock-9704/hardware. © Ground Control | the mount's slot height (1.70 +/-0.05, the datum for the printed rails' 1.80) and the antenna in the assembly view |
| `meshes/` | `supreme_step.stl` and `rb9704_step.stl`: our tessellations of the two board STEP files | the only inputs the validation chain reads (`../validation/clash_check.py`, `../validation/build_and_check.sh`) and the board bodies drawn in the `.scad`'s assembly and exploded views |

Two files of the delivered package are not duplicated here because this repository already holds them byte for byte: the board STEP `RockBLOCK-9704-SMA-2A.step` is [`v2/vendor/rockblock/RockBLOCK 9704-SMA-2A.step`](../../../v2/vendor/rockblock/) (52.7 MB, sha256 `44ec669bd683b7ee4d98f88535e0d98bf4a09cf471c74ae74a776c67088a85ce`), and the mount drawing `RB9704SMA-MOUNT-DIMS-REV-A.pdf` is [`v2/vendor/rockblock/rb9704-sma-dims.pdf`](../../../v2/vendor/rockblock/rb9704-sma-dims.pdf) (sha256 `968d7d5205517335db7ac8bd39f1852639b4683c01079573b93dd23a5184f343`). The package's own README names all of them under "Sources".

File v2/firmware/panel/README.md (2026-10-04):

# MeshSat field kit V2: panel controller firmware (board C, U3 RP2040)

MESHSAT-1357, Layer 12. **Prototype firmware for an unbuilt kit: no board C exists, nothing here has run on hardware,
and the target build has not been compiled** (this host has no arm toolchain and no pico-sdk). What has run: the
portable core and its 64 host unit tests, compiled with the host gcc 12.2 under `-std=c11 -Wall -Wextra -Werror
-pedantic -Wshadow -Wconversion`, all passing, and the Python checks of `v2/ecad/tools/tests/test_fw_panel.py` that bind
the code to the netlists and the contract pages.

**Round 3 (3 October 2026, branch `fnd/fw-r3` from set 28's `de45a5b4`):** Layer 5's third round (record l5r2,
`v2/docs/records/l5r2/L5-PANEL-R3.md`) decided this firmware's findings F-04 to F-13 in the contract and adopted 33 of its 36
session choices (`PANEL.md` section 9a, `HW-FW-CONTRACT.md` section 3.8). The firmware now follows every decided value:
F-05 (no TX lamp floor), F-07 (two modules lost is MASTER WARN), F-11 (board D's power-up levels) and the declined S-19 changed
the code; the rest it already did. Each decided value is bound by `test_fw_panel.py`'s `t_contract_*` cases (section 2).

**Round 4 (3 October 2026, branch `fnd/fw-r4` from `dea639a4` with Layer 5's `fnd/l5r4` at `0b3c058c` merged):** Layer 5
decided F-14 (record l5r4, `v2/docs/records/l5r4/L5-R4-SLOT-FAULTS.md`): ONE slot-fault rule for a module lost at start-up
and one lost while running, in `PANEL.md` section 5 and FW-C05, kept across a controller reset (FW-C02, V-C05). The firmware
follows it (section 1, FW-C05; finding F-14 closed, section 5), bound by `t_contract_f14_one_slot_fault_rule`.

The contract this implements: `v2/docs/PANEL.md` (cited P s.n), `v2/docs/HW-FW-CONTRACT.md` rows FW-C01 to FW-C15
(and the FW-A, FW-K rows they lean on), `v2/docs/feasibility/ZEROIZE.md` sections 3.4 and 3.5 (ZER), the pins of board
C's generator `v2/ecad/tools/gen_sch_c.py` and netlist `v2/ecad/pcb-c-display-c8/out/pcb-c-display.net`, and the
expander bits of boards A, B and D's netlists.

| Path | What |
|---|---|
| `include/panel.h` | the core's types, constants (each citing its statement) and API |
| `include/hal.h` | the hardware layer: every GPIO (`HAL_PIN_LIST`) and expander bit (`HAL_EXP_BIT_LIST`), the I2C map, the HAL calls |
| `src/panel_core.c` | the state machines with a millisecond tick: controls, indicators, lighting, sounder, e-paper model, slots, display select, shutdown, shore inhibit, EMCON, hot stop, margin hold, the power controls in part, the boot order |
| `src/zeroize.c` | the wipe journal and the crypto-erase sequence (ZER 3.4) and the boot table (ZER 3.5) over injected operations |
| `src/expander.c` | the seven PCA9555: the boot writes (outputs before configuration), the LED drive rule, the EXP_INT service, the switched loads' bits |
| `src/bus_recover.c` | the kit bus recovery (FW-K04) |
| `src/sensors.c` | board B's TMP117 (FW-C13's fallback) and board C's VEML7700 (P s.8), read off the kit bus |
| `src/hal_host.c` | the host stub of hal.h |
| `src/hal_rp2040.c`, `src/main_rp2040.c` | the pico-sdk implementation and main loop (NOT BUILT) |
| `CMakeLists.txt` | the target build (pico-sdk 2.3.1), NOT RUN |
| `Makefile`, `tests/` | the host build and tests: `make -C v2/firmware/panel test` |

## 1. What the core implements

Pure logic: `panel_tick(p, now_ms, in, out)` reads a sample of the inputs and writes the wanted outputs. The kit bus,
the secure element, the flash journal and the e-paper's command layer are reached through `panel_ops_t`, so the tests
replace each with a fake (a PCA9555 register model, an ATECC608B that can fail, a NOR flash that can tear, a BUSY line).

- **P s.3**: debounce 30 ms on every switch; PI_SHDN_REQ active low, only ever pulled low by its output enable (FW-A10);
  PI_KILL push-pull low from the first instruction (FW-A11); GPIO21 and GPIO22 inputs only; RAIL_SENSE present above 1.25 V.
- **P s.4**: the LED drive rule (on = output driving 0, off = input, never a 1), the outputs enabled one by one after
  boot, every expander's output registers before its configuration (FW-A08), DEV_EN kept 1.
- **P s.5, FW-C01, FW-C02, FW-C05, FW-C06**: the boot order; the SLOT_EN levels read and adopted at boot (all driven
  low first when the toggle is closed or a wipe is pending); the heartbeat (alive while toggling, lost 3 s after the
  last edge); a flat heartbeat 60 s after the rail came up is a slot fault, power-cycled once with 5 s off, then left
  off until the operator acts; since round 4 (F-14, record l5r4, FW-C05) ONE rule for both cases: a supervised slot
  (SLOT_EN high, no shutdown, hot stop, shed or ZEROIZE asked of it) is shown lost at once (3 s without an edge, or flat
  60 s after its rail came up; `EV_SLOT_FAULT`, MASTER CAUT); at 60 s without an edge counted from the later of its rail
  coming up and its last edge it is power-cycled once (`slot_flat_60s`, its one retry, `EV_SLOT_CYCLE`), and the next time
  left off (`EV_SLOT_OFF`) until the operator acts (`panel_slot_operator_retry` for the touch UI and the bridge, or MAIN);
  coming back never re-arms the retry; each slot's spent retry and left-off state are kept in their own flash region beside
  the wipe journal (`src/slotstore.c`) across a watchdog, RUN or SWD reset and cleared by a power-on reset (`panel_init`);
  the slots raised one at a time; HDMI_SEL follows the bridge, else the lowest live slot,
  never a dark one (slot 1 = both low, slot 2 = SEL1 high, slot 3 = SEL2 high, read from `gen_sch_b.py:1342-1348`).
- **P s.5, FW-C03**: a MAIN tap (INT low at least 32 ms), the PI button's short press or the bridge's command starts the
  clean shutdown: PI_SHDN_REQ low 200 ms, the heartbeats awaited, then PI_KILL high and held; the PI button held 8 s is
  PI_KILL at once.
- **P s.6, FW-C07**: the hardware lines are never driven (the output structure has no field for TX_INHIBIT_n,
  EMCON_HW or ZEROIZE_HW; the HAL refuses an output on GPIO21); every EMCON edge is reported for the bridge's software
  holds, MASTER CAUT steady; the RockBLOCK's ENABLE request (B:U6 RB_SW_IEN) low on EMCON and raised after a release
  only once a fresh RB_STATUS read is low (P corrections (17)).
- **P s.8**: DAY 100 %, NIGHT 15 %, NVG 2 % with red and amber indicators only, BLACKOUT 0 with every LED and the
  sounder dark; the backlight figures for the bridge; the TX lamp follows the one dimmer, keyed or not (F-05, round 3: the
  first contract's 10 % floor is withdrawn and `panel_light_duty` no longer takes the TX lamp's state).
- **P s.9**: MASTER WARN and CAUT (flash unacknowledged, steady after ACK, a cleared condition forgets its ACK; one
  compute module lost is MASTER CAUT and two lost MASTER WARN, F-07, `panel_modules_lost`),
  SOS ACTIVE, the bearer LEDs, SHORE and CHARGING from the charger's bits, MSG, the PI ring's 0.5 Hz heartbeat, the
  battery bar, the lamp test of all seventeen; TEST short press, hold 2 s, hold 5 s for the QR; SOS closed 2 s and every
  SOS indication; ZEROIZE closed 5 s with the abort, complete and incomplete indications; the sounder patterns; the
  e-paper's page selection, refresh pacing, full refreshes, power and BUSY sequencing; the bridge's indicators held
  when the USB link drops.
- **P s.10, FW-C08**: SHORE_INHIBIT boot low, raised only for 'inputs off' or the water-on-floor isolation, refused
  for any other reason, and refused until the bridge has warned while the pack cannot discharge; held through a link
  loss.
- **FW-C04, ZER 3.4 and 3.5**: the step-0 alarm, the PENDING record, C0 and C1 before any retry, the verifications
  against the created key and the recorded one, at most 6 GenKey commands before the deadline D, DONE, the modules told
  once the timed phase ends (by D plus the last operation's unwind; ZER gives 1.504 s), the slots cut on their confirmation or at 3.0 s, step 7's ten creates per slot, the journal's
  torn record reading PENDING (I3), and the five rows of the boot table.
- **PANEL.md s.4 and s.5, FW-C03 (DRAFTED by record l8r2)**: the PI button read on U1 P1.3 (PI_BTN_n, low = pressed)
  at every EXP_INT and the once-a-second poll, behind `pi_btn_wired` (`HAL_PI_BUTTON_WIRED` 0 until board C is regenerated
  with l8r2's draft: as generated the pin is a floating spare and must never read as a press).
- **FW-C13, FW-C14**: HOT-R1's four states decoded from A:U27 P1.5 at every EXP_INT and a poll every second (with a
  command byte other than 00h after each read); H1's actions and release (the heat stage's module first, then FW-C09 C1's restore 5 K below
  releases the others: S-19 declined), H2's page then PI_KILL, the TMP117 fallback
  with the reduced mode and the outlets off, and the start-up read before any slot rises.
- **FW-C15**: the margin hold's two-reading trigger at 68.65 C plus the reference's offset, its actions on A:U27 and
  B:U6, the SOS queued and told, and the restore 5 K under after 30 minutes; H1 overrides it.
- **FW-C09 in part**: the round-8 fallback (the pack readings stopped 10 s: the reduced mode, both outlets off) and
  C1's first stage (+50 C inside air or +55 C on a cell, restore 5 K below).
- **FW-K04**: nine SCL pulses and a STOP on a held bus, run by the target loop after a failed transfer and reported.
- **The kit-bus sensors**: board B's TMP117 (FW-C13's fallback) once a conversion, and board C's VEML7700 for the
  bridge (P s.8), both from the makers' sheets held in `v2/vendor/` (`src/sensors.c`'s header).

## 2. Statement to test

Every host test (64), from `tests/test_list.h` (the Python wrapper checks that each runs and passes, and that this table
names each).

| Test | Statement |
|---|---|
| t_debounce_30ms | P s.3: debounce 30 ms on every switch input |
| t_lighting_modes | P s.8: DAY, NIGHT, NVG (red and amber only), BLACKOUT, backlight |
| t_tx_lamp_follows_duty | P s.8 (F-05): the TX lamp follows the duty, NVG 2 % keyed, dark in BLACKOUT |
| t_rail_sense | P s.3 GPIO26 and s.8: the rail present above 1.25 V |
| t_led_drive_rule | P s.4: on = output driving 0, off = input, never a 1 |
| t_led_boot_one_by_one | P s.4: the outputs enabled one by one after boot |
| t_warn_caut_semantics | P s.9: flashing unacknowledged, steady after ACK |
| t_bridge_hold_on_link_drop | P s.9: the last state held when the USB link drops |
| t_msg_cleared_by_ack | P s.9: MSG cleared by ACK |
| t_battery_bar | P s.9: the battery bar 5 s, the lowest flashing below 10 % |
| t_pi_ring_heartbeat | P s.9: the PI ring at 0.5 Hz while a slot's bridge runs |
| t_sounder_patterns | P s.9: chirp, the double chirp 50/100/50 ms (F-06), SOS pattern, muted in BLACKOUT |
| t_epd_refresh_rules | P s.9: refresh pacing, full refreshes, power between refreshes (F-08) |
| t_epd_busy_polled | P s.9: BUSY polled before every command |
| t_test_short_press_ack | P s.9: TEST short press = acknowledge |
| t_test_hold_lamp_test | P s.9: hold 2 s = lamp test (F-06) |
| t_test_qr_while_held | P s.9: hold 5 s within 60 s of a show QR request |
| t_sos_hold_2s | P s.9, FW-C10: SOS closed 2 s, flipping back cancels |
| t_sos_indications | P s.9: the SOS indications; FW-C10 |
| t_sos_emcon_queue | FW-C10, V-C10: queued under EMCON |
| t_pi_button_logic | P s.5, FW-C03: the PI button (F-01) |
| t_emcon_edges | FW-C07; P corrections (17) |
| t_never_drives_hardware_lines | P s.6, FW-C07, FW-A10 |
| t_zeroize_abort_inside_5s | P s.9, FW-C04: the abort |
| t_zeroize_commit_sequence | FW-C04, ZER 3.4 steps 0 to 8 |
| t_zeroize_confirm_cuts_early | ZER 3.4 step 6; FW-C04 |
| t_zeroize_retry_policy | ZER 3.4 step 3 and step 7; FW-C04 |
| t_zeroize_incomplete | P s.9, ZER 3.4 step 7; FW-C04 |
| t_zeroize_rearm_on_return | FW-C04: re-arm on the toggle's return |
| t_journal_torn_reads_pending | ZER I3; FW-C04 |
| t_zeroize_boot_table | ZER 3.5; FW-C01 step 3; FW-C04 |
| t_boot_order | FW-C01 |
| t_boot_slot_adopt | FW-C02 |
| t_exp_outputs_before_config | FW-A08, FW-C01 step 4, P s.5 |
| t_hb_lost_3s | FW-C05 |
| t_slot_fault_cycle | P s.5, FW-C05: lost at start-up, cycled once, then off until the operator acts |
| t_slot_lost_while_running_cycled_once | FW-C05 (F-14): lost while running, shown at 3 s, cycled 60 s after its last edge |
| t_slot_lost_again_after_cycle_left_off | FW-C05 (F-14): lost again after a good cycle, left off; the retry re-arms |
| t_slot_not_supervised_while_stopping | FW-C05 (F-14): no supervision while a stop is asked (the hot stop) |
| t_slot_off_kept_across_controller_reset | FW-C05, FW-C02 (F-14): left off across a watchdog, RUN or SWD reset |
| t_slot_record_cleared_by_power_on | FW-C05 (F-14): a power-on reset clears every slot's state |
| t_slot_store_torn_keeps_previous | FW-C05 (F-14, S-37): a torn slot record keeps the previous state, never a pending wipe |
| t_hdmi_select | FW-C06, P s.5 |
| t_shutdown_main_tap | FW-C03, FW-A10, FW-A12 |
| t_shore_inhibit | P s.10, FW-C08 |
| t_hotr1_decode | FW-C14 |
| t_hot_stop_h1 | FW-C13: H1 |
| t_hot_stop_h2 | FW-C13: H2 |
| t_hot_tmp117_fallback | FW-C13, FW-C14: the line held high |
| t_hot_boot_read | FW-C14: the start-up read |
| t_hotr1_bus_lost | FW-C14: a bus that stops answering is the detector lost, never a stale held low |
| t_boot_main_tap | FW-C03, FW-A12: a MAIN tap during the boot |
| t_hot_boot_held_slot | FW-C14: a slot held up at boot, the line at 5 Hz |
| t_no_raise_while_zeroize_armed | FW-C04, D-03: nothing newly raised while ZEROIZE is armed or wiping |
| t_switch_closed_at_power_up | P s.9, FW-C10: SOS closed at power-up |
| t_tmp117_read | FW-C13, FW-C14: board B's TMP117 read off the bus, once a conversion |
| t_veml7700_read | P s.8: the VEML7700 reading for the bridge |
| t_se_absent_retried | FW-C04, ZER 3.5: the absent SE retried |
| t_margin_hold | FW-C15 |
| t_power_fallback | FW-C09 in part |
| t_modules_lost_caut_then_warn | P s.9 (F-07), CONOPS 4e: one module lost MASTER CAUT, two MASTER WARN |
| t_after_h1_restore_5k_below | FW-C13, FW-C09 (S-19 declined): the heat stage's module first, then C1's restore |
| t_pi_button_on_u1_p13_when_wired | P s.4 and s.5, FW-C03 (DRAFTED): PI_BTN_n on U1 P1.3, read only when wired |
| t_bus_recover | FW-K04, V-K02 |

The Python checks (`run.py fw_panel`): the host tests build and pass; every FW-C row is covered (section 3); hal.h's
30 GPIOs match U3's pins on board C's netlist (through `gen_sch_c.py`'s RP2040 table, read with `ast`); every expander
bit hal.h names matches its PCA9555 pin on boards A, B, C and D, and every address matches its A0 to A2 straps; the PI
button reaches no controller pin (F-01's evidence, which fails the day it is wired); no controller pin reaches the
panel LDO's enable (FW-C11); the e-paper messages quoted by P s.9, FW-C13 and FW-C15 are carried verbatim; 29 timing and
threshold constants equal the contract's figures, each with the words that must still stand in its page; the target
build keeps FW-C01's two rules and FW-C02's reset scope; and, since rounds 3 and 4, ten `t_contract_*` cases (F-04, F-05,
F-06, F-07, F-08, F-10, F-11, F-12, F-13, and F-14's FW-C05 rule: 3 s, 60 s from the later of the rail and the last edge,
rail off 5 s, one retry, kept across a controller reset, cleared by a power-on reset, re-armed by the operator) that read each decided value from the contract's own sentence and compare it with
what the core does, measured by the host program `tests/contract_probe.c` (`make -C v2/firmware/panel probe`): a contract row
the code contradicts fails by its finding's name, and a sentence that no longer parses fails as a contract change to re-read.

## 3. The FW-C rows

Machine-checked: every FW-C row of the contract is here; IMPLEMENTED and PARTLY rows are cited by a host test; the
other two statuses are cited by none.

| Row | Status | What the firmware does | What is owed |
|---|---|---|---|
| FW-C01 | PARTLY | steps 1 to 4 and 6 (`panel_init`, `boot_step`, `panel_exp_boot`); the E5 fix off and the BOOTSEL mask in `CMakeLists.txt` and `hal_reboot_to_bootsel` | step 5, the charger's registers (FW-A01 to A03, A16 to A18): no charger driver here |
| FW-C02 | PARTLY | the held levels read and adopted, all low first with a wipe due; a slot left off stays off across the reset (F-14); the watchdog with SIO, IO_BANK0 and PADS_BANK0 out of its scope and the SDK's early resets overridden (F-03); no ROM bootloader while a slot runs; the reset reason read | the boot reason reported (protocol, F-02); every hardware behaviour (V-C02) |
| FW-C03 | IMPLEMENTED | the MAIN tap, the PI short press and 8 s hold, the bridge's commands; the drafted PI input on U1 P1.3 read behind `pi_btn_wired` | the PI button's input is not wired on board C as generated (F-01; drafted by record l8r2, PROVISIONAL) |
| FW-C04 | PARTLY | the level-sensitive trigger, the abort, ZER 3.4's sequence and bounds, the journal, the boot table, the re-arm, an absent SE retried every 60 s, no slot newly raised while armed or wiping | the ATECC608B command layer (CryptoAuthLib and the bounded six-function HAL), P_A0 and P_B0 at enrolment, the modules told over the protocol (F-02); Z-EXP-A to C |
| FW-C05 | IMPLEMENTED | inputs without pad pulls, alive while toggling, lost after 3 s, the display re-elected; the one slot-fault rule of F-14 (round 4): shown at the loss, cycled once at 60 s from the later of the rail and the last edge, then left off until the operator acts, the state kept across a controller reset and cleared by a power-on reset | the e-paper's naming of the slot (the rendering, section 4); a bridge message that suspends supervision for a planned restart (MESHSAT-837) |
| FW-C06 | IMPLEMENTED | follow the bridge, else the lowest live slot, never a dark slot | |
| FW-C07 | IMPLEMENTED | GPIO21 an input only, every EMCON edge reported, MASTER CAUT steady, EMCON on the e-paper (its own page, and in the SOS pages) | the software holds themselves (queue, AT+CFUN, rfkill) are the bridge's |
| FW-C08 | IMPLEMENTED | boot low, only the two reasons, the warning first, never a charge hold | |
| FW-C09 | PARTLY | the round-8 10 s fallback, C1's first stage and its restore 5 K below (which also releases the slots held after H1) | C1's second stage ("reached again there"), C2, C3, C4 and K1 to K5 (`POWER-THERMAL.md` 7.2, PROVISIONAL, not read into this firmware); the readings reach the panel only over the protocol (F-02) |
| FW-C10 | IMPLEMENTED | the 2 s hold, the indications, queued under EMCON, the cancel | the sending is the bridge's |
| FW-C11 | NOT THE FIRMWARE'S | no controller pin reaches U5's EN (on +5V): the firmware has no means to switch its 3.3 V (`t_panel_3v3_cannot_be_switched_by_firmware`) | |
| FW-C12 | OWED | nothing: the wire format (MESHSAT-837) is defined nowhere (F-02); `panel_bridge_t` is only the decoded content the core reads, and the switch edges are queued as events | the wire format, the USB composite device (CDC and HID), the codec, V-C12 |
| FW-C13 | PARTLY | H1 and H2, the clean-shutdown request, the loads off on A:U27 and A:U28, each slot dropped once it has stopped, the release and the heat stage's one module (then FW-C09's restore, S-19 declined), the TMP117 fallback on board B's TMP117 read off the bus once a conversion | the CHRG_INHIBIT bit's write (FW-A19's charger driver; the core raises the flag); the hottest reading on the e-paper (the rendering, section 4) |
| FW-C14 | IMPLEMENTED | the four states, the start-up read, the slot found held up, the EXP_INT service with the command byte, the 1 s poll | |
| FW-C15 | PARTLY | the trigger, the actions on A:U27 and B:U6, the SOS queued and told, MASTER CAUT, the page, the restore, H1's precedence | the Geiger off (the sensor controller, over the protocol), the module idled (the bridge), the CHRG_INHIBIT write, the reference's offset (T-H1) |

## 4. Not implemented, and owed

- **The bridge protocol (FW-C12)**: finding F-02. Until it exists the core runs as if no host were present.
- **The e-paper's command layer and rendering**: the PDi E2370KS0C1's iTC sequence (UltraChip UC8253C class, sheet held
  as `v2/vendor/pdi/ultrachip-uc8253c-a0.6.pdf`), the fonts, the pages' fields and the QR encoder. The core decides
  which page, when, full or partial, and sequences EPD_PWR_n and BUSY; `panel_epd_ops_t.send` is a stub.
- **The charger (FW-A01 to A23)**: no register is written; the core raises the CHRG_INHIBIT flags (hot, margin) and
  reads the SHORE and CHARGING bits as inputs a driver would fill.
- **The secure element**: CryptoAuthLib is not vendored; on the target every SE call fails, so the boot takes "the SE
  does not answer" and a commit ends INCOMPLETE with the slots held off (fail secure).
- **The USB device**, and the kit bus segment buffer of FW-K05 (OWED in the contract). The VEML7700's lux per count at
  the chosen setting is INFERRED by scaling (sensors.c); Vishay's application note is not held.
- **The pico-sdk build**: never compiled; the SDK names were read from pico-sdk 2.3.1 (section 6).

## 5. Findings

Each is raised for the page or board named; nothing in a contract, record, generator or PANEL.md was edited.

| ID | Severity | Finding | Exact place | Owner | Round 3 (record l5r2, `L5-PANEL-R3.md`) |
|---|---|---|---|---|---|
| F-01 | major | The PI button reaches no controller pin. SW_PI's contacts (PIJ2_A, PIJ2_B) pass FB3 and FB4 to J_PIJ2's two lands (PIJ2_A2, PIJ2_B2) and to U11's clamps only: no U3 GPIO, no expander input, neither on GND, and no other board has a mating lead. PANEL.md s.5 and FW-C03 have the controller read it; ASSEMBLY.md says "the panel controller reads it; nothing leaves the backer"; the generator's own note says PIJ2_A2 is the LTC2954's INT on board A. Every one of the 30 GPIOs is used; the expanders' spares are free (U1 P1.3 to P1.7, U2 P1.1 to P1.7). The firmware's logic is done and tested on an input the target HAL cannot fill (`HAL_PI_BUTTON_WIRED 0`) | `gen_sch_c.py:324-326`, `:333`; netlist nets /PIJ2_A2 and /PIJ2_B2; `ASSEMBLY.md:127`; `PANEL.md:149` | board C's author | drafted by record l8r2 (U1 P1.3, PI_BTN_n), PROVISIONAL until board C is regenerated; the code reads it behind `pi_btn_wired` (`t_pi_button_on_u1_p13_when_wired`); `t_pi_button_reaches_no_controller_pin` fails the day the netlist wires it, to flip `HAL_PI_BUTTON_WIRED` |
| F-02 | major | The bridge protocol's wire format (MESHSAT-837) is defined nowhere: not in the meshsat repository (docs, internal, proto, and no commit message names MESHSAT-837), not in the HAL repository, not in this tree, and the YouTrack issue carries a goal, no format. Nothing of it is implemented. Consequence on the target: no bridge input (the SOS "NO HOST" indication, the bridge's LEDs dark, every switched load off, SHORE_INHIBIT never raised), no pack readings (FW-C09, FW-C15's reference, the battery bar), and ZER 3.4 step 5 has no channel, so step 6 waits for the 3.0 s alarm | `PANEL.md:215`; `HW-FW-CONTRACT.md:461` | MESHSAT-837's owner | open (MESHSAT-837); round 3 names the bridge protocol as the operator's retry path (F-09) |
| F-03 | major | FW-C02's reset scope cannot keep SLOT_EN by itself: pico-sdk 2.3.1's `runtime_init_early_resets()` resets IO_BANK0 and PADS_BANK0 on every boot (`runtime_init.c:56-70`), so the firmware overrides that weak function. Whether the PSM's RESETS bit must also be cleared is INFERRED (`hal_watchdog_start`), for V-C02. And ZER 3.4 step 0's backstop ("SLOT_EN1..3 return to inputs" on a watchdog reset) no longer holds under FW-C02: a hang during a wipe is cut by the reset and then the boot path, which drives every SLOT_EN low first with the toggle closed or a PENDING record, at the watchdog period (1 s here) plus the boot's first instructions | `HW-FW-CONTRACT.md` FW-C02; `feasibility/ZEROIZE.md:259-264` | the contract's writer; ZEROIZE.md's owner | carried into FW-C02 by `HW-FW-CONTRACT.md` 3.8 as the firmware's finding; the PSM bit read at V-C02 |
| F-04 | minor | PANEL.md s.4 orders board C's boot as "first writes the configuration registers so every LED bit is an input, then the output registers to 0"; s.5 and FW-A08 order every expander's output registers first. Both are safe on U1 and U2 (every bit written 0, off is an input); the firmware writes outputs first everywhere, then configuration all inputs, then the outputs one by one | `PANEL.md:139` against `PANEL.md:147` | PANEL.md's writer | decided: outputs before every configuration write (PANEL.md 4, FW-A08, S-10); the code already did; `t_contract_f04` |
| F-05 | minor | NVG's 2 % and "the TX lamp is never dimmed below 10 % duty" share one rail (LED_RAIL behind Q1). The firmware raises the whole panel to 10 % while TR_APRS reads keyed or the lamp test lights the TX lamp, so in NVG the lit red and amber LEDs rise to 10 % for a key-down | `PANEL.md:192`, `:195` | PANEL.md's writer | decided: the floor withdrawn, the TX lamp follows the duty; CODE CHANGED: `panel_light_duty` (no TX argument) and `panel_tick`; `t_contract_f05` |
| F-06 | minor | The lamp test's sound: "a chirp" in the controls, "double chirp (lamp test)" in the sounder patterns. Taken: the double chirp | `PANEL.md:201`, `:209` | PANEL.md's writer | decided: the double chirp 50/100/50 ms (S-15); the code already did, now named `PANEL_DCHIRP_*`; `t_contract_f06` |
| F-07 | minor | A slot fault is in both MASTER WARN's red list and MASTER CAUT's amber list; s.5 names MASTER CAUT. Taken: MASTER CAUT | `PANEL.md:199`, `:147` | PANEL.md's writer | decided: one slot fault MASTER CAUT, two modules lost MASTER WARN (CONOPS 4e); CODE CHANGED: `panel_modules_lost`, `indicators`; `t_contract_f07` |
| F-08 | minor | "Refresh at most once a minute" would delay the QR's removal (the glass keeps it with the power off), the SOS and the ZEROIZE pages. Taken: a change of page refreshes at once; the minute bounds the idle page's content | `PANEL.md:203` | PANEL.md's writer | decided as the firmware did; PDi's least interval owed to Layer 6 (L5R3-F03); `t_contract_f08` |
| F-09 | minor | "Until the operator acts" names no control. The core offers `panel_slot_operator_retry()` for the bridge (owed, F-02); no panel control does it | `PANEL.md:147` | PANEL.md's writer | decided: the retry over the bridge protocol (owed, F-02) or a restart with MAIN, after which every slot is raised again (the code keeps no fault across a restart) |
| F-10 | minor | At start-up FW-C14 says a 5 Hz line raises no slot "until it is back at 1 Hz"; FW-C13 leaves H1 only after 1 Hz AND 30 minutes. The firmware enters H1 at boot and waits for both (the stricter) | `HW-FW-CONTRACT.md` FW-C13, FW-C14 | the contract's writer | decided: the stricter rule (H1 dated at boot, 1 Hz and 30 minutes); the code already did; `t_contract_f10` |
| F-11 | minor | Board D's U16 outputs X_SA_PD, X_AMP_EN and X_MMUTE (FW-D01) have no stated boot level; the firmware writes 0 (S-11), which may hold the SA868 powered down until the bridge acts | `HW-FW-CONTRACT.md` FW-D01; `gen_sch_d.py:930` | board D's author | decided: X_SA_PD 1, X_AMP_EN 1, X_MMUTE 0, the generator's levels; S-11 declined; CODE CHANGED: `EXP_BOOT` (0x60, configuration 0x1F); `t_contract_f11` |
| F-12 | minor | FW-C15's "an SOS raised meanwhile is queued as under EMCON and the operator told" gives no message; the EMCON message ("OPEN EMCON TO SEND") would be wrong. Taken: "SOS QUEUED: MARGIN HOLD, COOLING" | `HW-FW-CONTRACT.md` FW-C15 | the contract's writer | decided: the firmware's text, in PANEL.md 9 and FW-C15; `t_contract_f12` |
| F-13 | observation | HDMI_SEL's encoding is in no contract page; read from board B: slot 1 both low, slot 2 SEL1 high, slot 3 SEL2 high (U3 and U4 cascade, U519 and U520 enables) | `gen_sch_b.py:1342-1348` | PANEL.md's writer | decided: the encoding as read; the code already did, now `panel_hdmi_encode`; `t_contract_f13` |
| F-14 | minor | A compute module lost while running: `CONOPS.md` section 4e's row "a compute module lost" handles it as "the slot is cycled once and then left off until the operator acts (`PANEL.md` section 5)", but PANEL.md section 5's trigger is a heartbeat flat for 60 s after the rail came up, the start-up case. The firmware follows PANEL.md 5's trigger: a module that stops while running is shown lost (MASTER CAUT, two lost MASTER WARN, F-07) and is not power-cycled | `CONOPS.md` section 4e's fault table; `PANEL.md` section 5 | Layer 5 (PANEL.md's writer) | CLOSED by Layer 5 round 4 (record l5r4): one rule for both cases in PANEL.md 5 and FW-C05, CONOPS 4e governing; the firmware follows it in round 4 (`slots_policy`, `slot_flat_60s`, `src/slotstore.c`, `panel_init`); `t_contract_f14_one_slot_fault_rule` |
| F-15 | minor | FW-C05 clears the slot state on a power-on reset named as "CHIP_RESET HAD_POR", and record l5r4's list says "after a watchdog, RUN or SWD reset (`HAD_POR` clear)". The RP2040 datasheet says CHIP_RESET gives "the source of the most recent chip-level reset" (2.12.7), and a watchdog reset is not chip-level, so HAD_POR still reads 1 after a watchdog reset that follows a power-on; on HAD_POR alone a watchdog reset would clear a slot left off. The firmware takes a power-on reset as HAD_POR with the watchdog's REASON zero ("Both bits are zero for the case of a hardware reset", 4.7, Table 548): `hal_reset_was_power_on` | `HW-FW-CONTRACT.md` FW-C05; `records/l5r4/L5-R4-SLOT-FAULTS.md` section 7 item 4; `v2/vendor/rp2040/rpi-rp2040-datasheet.pdf` 2.12.7 and 4.7 | Layer 5 (the contract's writer) | raised in round 4 (`fnd/fw-r4`); the code follows the datasheet, V-C05's watchdog reset checks it |

## 6. Session choices

Taken by the session under the owner's standing rule of 26 September 2026 where the contract leaves the firmware a
choice. Each is reversed by changing the named constant or line.

| ID | Choice | Why | Reverse | Contract (round 3) |
|---|---|---|---|---|
| S-01 | hold times run from the debounced edge | never shorter than stated | `controls_*` | adopted (PANEL.md 9a) |
| S-02 | MASTER WARN and CAUT flash at 4 Hz; the low battery LED at 2 Hz | inside P s.9's 3 to 5 Hz | `PANEL_FLASH_*` | adopted (PANEL.md 9a) |
| S-03 | the slots raised 1 s apart | "one at a time" with no interval | `PANEL_SLOT_STAGGER_MS` | adopted (PANEL.md 9a; FW-C01 in 3.8) |
| S-04 | the operator's retry is a call for the bridge | F-09 | `panel_slot_operator_retry` | adopted (PANEL.md 9a; F-09) |
| S-05 | a clean shutdown waits at most 60 s for the heartbeats | FW-C13's figure; FW-C03 gives none | `PANEL_SHDN_WAIT_MS` | adopted (FW-C03 in 3.8) |
| S-06 | "no host" = no bridge session | the panel cannot tell a module without its bridge from no module | `page_select`, `indicators` | adopted (PANEL.md 9a) |
| S-07 | HOT-R1: five or more edges in 2 s = 5 Hz, a held line after 3 s, 1 Hz only after 2 s of samples; polled every 50 ms during the start-up read | FW-E10 sends one edge a second at 1 Hz and five at 5 Hz | `panel_hot_classify` | adopted (FW-C14 in 3.8) |
| S-08 | H2 drives PI_KILL once its page is shown or after 30 s | the page first, as FW-C13 orders | `PANEL_H2_PAGE_WAIT_MS` | adopted (FW-C13 in 3.8) |
| S-09 | the watchdog's period 1 s | over the 235 ms worst GenKey; ZER leaves it TBD | `PANEL_WATCHDOG_MS` | adopted (FW-C02 in 3.8) |
| S-10 | every configuration write preceded by an output write of 0 | an expander reset by a brownout returns to FFh | `expander.c` | adopted (FW-A08 in 3.8; F-04) |
| S-11 | board D's U16 outputs written 0 | F-11 | `EXP_BOOT` | NOT ADOPTED: it would hold the SA868 powered down; FW-D01 takes the generator's power-up levels (F-11). The code now writes X_SA_PD 1, X_AMP_EN 1, X_MMUTE 0 |
| S-12 | the texts the contract does not quote: IDLE, ENROLMENT QR, SOS SENT, the SE's absence, the margin hold's SOS, EMCON ON | none stated | `panel_page_text` | adopted in part: the margin hold's text (F-12, PANEL.md 9 and FW-C15); the other texts stay the firmware's wording |
| S-13 | both LIGHTING inputs low (not possible on a sound toggle) = the dimmer lit mode, flagged | fail dim | `panel_light_mode` | adopted (PANEL.md 8 and 9a) |
| S-14 | battery LED k lit above 20(k-1) % | no empty bar from 10 to 19 % | `indicators` | adopted (PANEL.md 9a) |
| S-15 | the double chirp 50 on, 100 off, 50 on; the incomplete pulses 200 apart | none stated | `sound_level` | adopted (PANEL.md 9; F-06) |
| S-16 | a page change refreshes at once | F-08 | `epd_step` | adopted (PANEL.md 9; F-08) |
| S-17 | HOT-R1 unreadable at start-up = held high (the detector lost) | fail to the TMP117 fallback | `boot_step` | adopted (FW-C14 in 3.8) |
| S-18 | a 5 Hz line at start-up enters H1 with the stop at boot | F-10 | `boot_step`, `hot_step` | adopted (FW-C14 in 3.8; F-10) |
| S-19 | after H1 only the heat stage's module (slot 2 as board B is generated) runs until the next start | FW-C09's restore is not implemented | `heat_stage_only` | NOT ADOPTED: the firmware's interim while FW-C09's restore was unimplemented; the contract's restore 5 K below stands. The code now raises the heat stage's module first and lifts the limit once it runs and C1's restore condition holds (`power_controls_step`); with no pack readings (no bridge, F-02) the restore cannot be judged and the limit stays |
| S-20 | the margin reference's offset 0 until T-H1 calibrates it | FW-C15 PROVISIONAL | `PANEL_MARGIN_REF_OFFSET_MC` | adopted (FW-C15 in 3.8) |
| S-21 | after a complete wipe the slots power again when the toggle returns | ZER 3.5's re-armed row | `controls_zeroize` | adopted (PANEL.md 9a; FW-C04 in 3.8) |
| S-22 | the lamp test fires at 2 s on the way to a 5 s QR hold | both statements are unconditional | `controls_test` | adopted (PANEL.md 9a) |
| S-23 | NVG's red-and-amber rule applies to the lamp test | light discipline | `panel_tick` | adopted (PANEL.md 9a) |
| S-24 | the sounder sounds in DAY, NIGHT and NVG; ACK mutes the SOS and incomplete patterns until the condition rises again | P s.8 mutes only BLACKOUT | `sound_level` | adopted (PANEL.md 9a) |
| S-25 | ZEROIZE arming and incomplete force MASTER WARN to flash, complete forces it steady, whatever the ACK | P s.9's ZEROIZE indications are specific | `indicators` | adopted (PANEL.md 9a) |
| S-26 | the pack fallback only after the readings were seen once | a bridge not yet booted is not a lost sensor controller | `power_controls_step` | adopted (FW-C09 in 3.8) |
| S-27 | with no bridge every switched load stays off | the loads' policy is the bridge's | `panel_exp_write_kit` | adopted (FW-C09 in 3.8) |
| S-28 | the EXP_INT service reads every input expander and writes the command byte to each | FW-C14 names U27; harmless on the others | `panel_exp_service` | adopted (FW-C14 in 3.8) |
| S-29 | this controller's own pull on PI_SHDN_REQ, and 5 ms after it, is never read as a MAIN tap | the line is one wired-OR net | `PANEL_OWN_PULL_GUARD_MS` | adopted (FW-C03 in 3.8) |
| S-30 | an EXP_INT held low is serviced at most every 5 ms; a failed LED write retried after 100 ms | a dead target must not stall the loop at 10 ms a transfer | `PANEL_EXP_INT_MIN_MS`, `PANEL_LED_RETRY_MS` | not a contract value (internal to the firmware, PANEL.md 9a); kept as the firmware's internal interval |
| S-31 | with every slot dark the display selection stays where it was | no live slot to choose; board B's enables pass no picture from a dark slot | `display_select` | adopted (PANEL.md 5 and 9a; FW-C06 in 3.8) |
| S-32 | HOT-R1 decided only on reads at most 1.5 s old; 1.5 to 3 s without a read keeps the last verdict; over 3 s is the detector lost | a dead bus must not age a stale low into H2 and kill the kit | `panel_hot_classify` | adopted (FW-C14 in 3.8) |
| S-33 | a TEST, SOS or PI switch already closed at power-up counts its hold from the controller's start (an SOS toggle left closed arms SOS 2 s after boot) | the toggles are maintained; a hold cannot be shorter than stated | `sample_switches` | adopted (PANEL.md 9a) |
| S-34 | no slot is newly raised while ZEROIZE is armed (the 5 s) or wiping; a running slot is left to step 6 | fail secure: D-03 cuts the slots | `zeroize_blocks_raise` | adopted (PANEL.md 9a; FW-C04 in 3.8) |
| S-35 | an absent secure element is retried every 60 s (two GenKey-public reads, about 0.26 s of the loop); its answer clears the warning | ZER 3.5 says it is retried and states no period | `PANEL_SE_PROBE_MS` | adopted (FW-C04 in 3.8) |
| S-36 | the TMP117 polled every 250 ms and counted once per Data_Ready (its reset setting converts each second); the VEML7700 at gain x1/8 and 100 ms (to about 35 klx), polled each second | "two readings in a row" are two conversions; daylight without saturation at NIGHT's cost of 0.54 lx steps | `PANEL_TMP117_POLL_MS`, `sensors.c` | adopted in part: the definition of a reading (FW-C13 in 3.8); the polling period and the VEML7700's gain stay internal |
| S-37 | each slot's spent retry and left-off state kept in a flash sector of its own beside the wipe journal, append-only, the last valid record winning and a torn one skipped | FW-C05 asks for it "with the wipe-pending record"; inside the journal ZEROIZE.md's invariant I3 would read a slot record torn by a power loss as a pending wipe and crypto-erase the keys | `src/slotstore.c`, `SLOTSTORE_OFF` | new in round 4; the contract's "with the wipe-pending record" read as beside it, in the same flash |

## 7. What needs the hardware

Bring-up of board C, in this order: power with the ribbon out and SWD on TP1 to TP3; the first target build (section 8);
the pins (each GPIO's level against hal.h); the expanders at 0x22 and 0x23 and the LED rule (a ghosted LED means a 1
was driven); the kit bus at 100 kHz on the scope (V-K01); then the ribbon in. The verification rows this firmware
feeds, none run: **V-C01** (no glitch on any enable but DEV_EN, the slots only after ZEROIZE_SW), **V-C02** (watchdog,
RUN and SWD resets with three slots running; F-03's INFERRED PSM bit), **V-C03** (MAIN tap, PI short and 8 s, the
force-off), **V-C04**, **V-C05** (a bridge stopped: lost within 3 s, the display moved), **V-C08**, **V-C09**, **V-C10**,
**V-C12** (after F-02), **V-C13** (P15 and E3-H), **V-C15**, **V-K01** to **V-K03**, **Z-EXP-A** to **Z-EXP-C** (the
secure element), **E-01** to **E-12** (EMCON), and the e-paper's first refresh (BUSY, the boost).

## 8. Building

Host tests (any host with gcc and make; nothing is written into the tree with `BUILD=` elsewhere):

    make -C v2/firmware/panel test
    env -C v2/ecad/tools/tests python3 run.py fw_panel

Target (owed; not run here): pico-sdk 2.3.1, arm-none-eabi-gcc, CMake 3.13 or later:

    export PICO_SDK_PATH=/path/to/pico-sdk   # tag 2.3.1
    cmake -S v2/firmware/panel -B build-rp2040 && cmake --build build-rp2040   # meshsat_panel.uf2 / .elf

Flash by SWD (TP1 SWCLK, TP2 SWDIO, TP3 RUN), never through the ROM bootloader while a slot runs (FW-C02).

The pico-sdk names `hal_rp2040.c` and `CMakeLists.txt` use were read from pico-sdk 2.3.1 on 3 October 2026
(`https://raw.githubusercontent.com/raspberrypi/pico-sdk/2.3.1/src/...`, BSD-3-Clause, consulted, not filed), sha256
first 16 hex: `rp2_common/pico_runtime_init/runtime_init.c` 7246c432e8b91c87, `rp2_common/hardware_watchdog/watchdog.c`
e7052da8894a7f12, `rp2040/hardware_regs/include/hardware/regs/psm.h` 99db9c7f82033171, `.../regs/resets.h`
bc261dcd8268c225, `.../regs/vreg_and_chip_reset.h` 002454b252fece95, `.../regs/intctrl.h` 76d1205144a953c7,
`rp2040/hardware_structs/include/hardware/structs/timer.h` 9325fe9694d9d6c8, `rp2_common/hardware_irq/include/hardware/irq.h`
85fabc3046de2b00, `rp2_common/hardware_resets/include/hardware/resets.h` 3688d3a282705b79,
`rp2_common/pico_bootrom/include/pico/bootrom.h` df34abac2ede9284, `common/pico_time/include/pico/time.h`
5cb0f594effa694e, `rp2_common/hardware_timer/include/hardware/timer.h` 5498220e5310d49e, `rp2_common/hardware_i2c/include/hardware/i2c.h`
ba330ff219f3844a, `rp2_common/hardware_flash/include/hardware/flash.h` 34bcc266f4535e6c, `rp2_common/tinyusb/CMakeLists.txt`
293d51840416b722.

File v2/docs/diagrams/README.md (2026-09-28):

# Diagrams of the V2 field kit (handover layer 4)

MESHSAT-1357, 27 September 2026. **Every diagram here is a design diagram of an unbuilt prototype.** No V2 board has
been fabricated, ordered or powered, no kit has been built, fitted to a case or field deployed, and nothing drawn here
has been measured. Each rendered file says so in its own title or footer.

**Status: rebuilt at `2781cee6` (29 September 2026, integration set 9's line, MESHSAT-1357), all 11 diagrams.** The
rebuild follows sets 6 to 9: the power tree types board D's feed as S-99 (decision 55) made it, VBAT to +5V_D8IN through
the TPS62933 buck U41 (enabled by RAIL_EN) and +5V_D8IN to +5V_D8 through the eFuse U23, where it had +5V_DEV to +5V_D8;
its sweep still accepts 15 substitutions, as before. The control lines follow board B's per-slot EMCON_HW gates (the
SN74LV1T08 map added to `tools/netlist.py` from TI SCLS739F Table 5-1, which the build refused without). Rendered on the
rented box (Mermaid CLI 11.12.0, Node 18, matplotlib 3.6.3); `build.py --check` reads 11 of 11 current against
`MANIFEST.json`; the readback (`readback.py`, its output in `v2/docs/records/diag/readback.log`) reports no problem: every
SVG parses, carries no foreignObject and states that it is a design diagram of an unbuilt prototype, and every PDF
prints at its drawing's natural size. The paragraph below is the record of the build at `b7f96784`.

**Status: drawn at `b7f96784`, with round 8 on all six boards and set 5 on boards A, B, D and E.** The r8int5 integration
(27 September 2026, branch `fnd/r8int5`) rebuilt every diagram again from the tree at `b7f96784` (netlists A `da05dc02bc1e612f`, B
`8b78c59754a6a0c7`, C `11eabc2dddca5161`, D `76700a687eb6187f`, E `d6137f50059e5cbc`, P `085f833362fbbda8`; `pcb_energy_chain.yaml` `a09ca0293afd1f7c`), after set 5 changed
the netlists of A, B, D and E. `power_tree.py` refused them as stream w3g left it, and follows them now: board E's
tracker stage names Q3, U5 and Q6 (R5 senses in the bottom switches' leg since S-47, off the PV_P to TRK_OUT path),
the VIN_RAW lead runs from board E's P_VR to board A's J_VR1 to J_VR4 (EQ-16), and the legend calls board B's
coin-cell net VBAT_RTC (W3B-R1). The case drawings now read r8int4's case release (`c351115d`). The rest of this page
is stream w3g's record of its rebuild at `38dcd764`, with the counts and findings of `b7f96784` given where they differ.
`build.py --check` reads 11 of 11 current against `MANIFEST.json`, whose `tree` is `b7f96784`.

Stream w3g's rebuild: every diagram was rebuilt on 27 September 2026 from
the tree at `38dcd764` (netlists A `3a786cf31614fe63`, B `adcc3c6736c90e9f`, C `11eabc2dddca5161`, D
`0dad82b4b6a79290`, E `f3c1ad6153002976`, P `085f833362fbbda8`; `pcb_energy_chain.yaml` `97c6afce242a590b`), each
netlist's sha256/16 in its own board box, with this folder's tools and the `ARCHITECTURE.md` reference lines of the
same rebuild. `python3 v2/docs/diagrams/tools/build.py --check` reads 11 of 11 current against `MANIFEST.json`, whose
`tree` is `38dcd764` and whose `inputs_differing_from_the_tree` names exactly the files this rebuild changed
(`ARCHITECTURE.md` and the tools); once they are committed as they stand, the check stays at 11 of 11 until an input
moves. The drawings made at `e3aedb25`, before round 8, are replaced: round 8 put board D's transmit chain behind a
load switch (`+5V_TX`, U21), split board B's EMCON line per slot (`EMCON_ON1..3`) and replaced the gates on the EMCON
lines of boards A, B and C, and the power tree and the control lines now show that.

The editable originals stay where they are: the Mermaid blocks in `v2/docs/ARCHITECTURE.md` and in the battery review
packet, the netlists under `v2/ecad/pcb-*/out/`, and the geometry sources named below. This folder holds readable
renderings of them, the tools that make them, and `MANIFEST.json`, which ties every rendered file to the sha256/16 of
each input it was made from.

## What is here

| Diagram | Shows | Drawn from | Does not show |
|---|---|---|---|
| `svg/arch-2-context.svg` | the kit in its context: operator, local networks, bearers, power inputs | `ARCHITECTURE.md` section 2 (its Mermaid block, unchanged) | anything the page's own block does not |
| `svg/arch-3-2-board-interconnect.svg` | the seven boards and the contracts between them | `ARCHITECTURE.md` section 3.2 | pin maps (they are in `pcb_interfaces.yaml`) |
| `svg/arch-4-1-power-tree.svg` | the power tree as the page summarises it | `ARCHITECTURE.md` section 4.1 | the netlist check of each stage (see `power-tree` below) |
| `svg/arch-4-3-power-up.svg` | power-up states S0 to S5 | `ARCHITECTURE.md` section 4.3 | timing; the SLOT_EN hold, which is in no generator |
| `svg/arch-5-5-lanes-and-fabric.svg` | PCIe, USB banks, Ethernet and display per slot | `ARCHITECTURE.md` section 5.5 | the supervisors and their CAN fabrics; channel budgets (FB-FAB-7) |
| `svg/battery-protection-states.svg` | the pack's protection states | `review-packets/battery/PROTECTION-ARCHITECTURE.md` section 4 | thresholds (in `PRIMARY-CONFIGURATION.md`) |
| `svg/battery-charger-states.svg` | the charger's state sequence with its host present or silent | `review-packets/battery/CHARGER-STATE-SEQUENCE.md` (the block sits under its section 7 heading, which the title quotes) | bench results (FW-A15 is open) |
| `svg/control-lines.svg` | TX_INHIBIT_n, EMCON_HW, board B's per-slot EMCON_ON1..3, ZEROIZE_SW, ZEROIZE_HW, SLOT_EN1..3, PI_KILL and SHORE_INHIBIT across boards C, B, A, D and E: the part driving each line and every part it reaches, followed through logic gates (pin maps from the makers' sheets, `netlist.py`), FET gates and series resistors, with the pulls, filters and connector pins | the committed netlists, read by `tools/control_lines.py`; pins checked at both ends and against `v2/ecad/tools/pcb_interfaces.yaml` | direction as firmware sets it, timing, test points (listed in `control-lines.md`), PI_SHDN_REQ, HDMI selects, heartbeats, the kit I2C bus, the SLOT_EN hold (in no generator); whether a line's state is proved (`feasibility/EMCON.md`) |
| `svg/power-tree.svg` | board P's cells to every rail on boards E, A, B, C and D, the three inputs, the leads between boards, the loads that leave the boards; board D's `+5V_TX` behind U21; the stages of `pcb_energy_chain.yaml` in red with their declared currents | the committed netlists and `v2/ecad/tools/pcb_energy_chain.yaml`, read by `tools/power_tree.py`; which parts make each stage is typed in the tool and checked against the netlist on every build (method and limits in `power-tree.md`) | currents drawn, losses, heat, which rail is on in which power state, grounds and returns, clamps, the CM5 modules' own rails |
| `svg/case-plan.svg` | the Peli 1450 cavity, the 1450PF window, face plate C1, the setting legs C6, boards A, B, C (backer strips), D, E, E5, the 4S3P block and board P, the rods, the blind-mate row, the arrestors of C2 and the connector plate of C3; the superseded as-coded plate and wall jacks in grey | `v2/vendor/peli/frame_seat.py` and its output, `v2/vendor/peli/case_margins.py`, `v2/ecad/tools/panel1450.py`, the board generators' constants, `pcb_board_facts.yaml` (checked) | parts on the boards, cables, the pack's hold-down (not designed, S-27), the lid, tolerance bands; board P's position is INFERRED |
| `svg/case-zstack.svg` | the same arrangement in Z along X: floor, walls, rim, shoulder, rib tops, every board, the CM5 heatsinks, the pack block, the legs, the 1450PF frame in section (ring on the leg pads, skirt down to its bottom 86.00, outer face, gasket step and flange), the face plate with its range, the Xenarc body and margin M1, the arrestor axis; the as-coded face top and jacks in grey; detail A enlarges the frame at the end wall with M20 and M21d | as above, plus `v2/cad/render/scene.py` for the heights of E5, A and D | the backer ring, the e-paper, the PA under the plate, cables, the lid tray, tolerance stacks, the frame's corner arcs, insert bores and gasket, what the pack block stands on (S-27) |

Each diagram has a PDF copy in `pdf/`, printed at the drawing's natural size (the wide ones are large-format pages:
the power tree 6360 x 1476 pt, the control lines 4940 x 1202 pt; zoom to fit or print in tiles). The Mermaid sources
the SVGs were rendered from are in `src/`: the seven copied out of the documents carry only an added title (document,
section, line range and the document's sha256/16; the tree revision is in `MANIFEST.json`, since a file cannot name
the commit that contains it); `control-lines.mmd` and `power-tree.mmd` are generated. The netlist readings behind the
generated diagrams are in `control-lines.md` and `power-tree.md`, and every number of the case drawings with its
source is in `case-drawings.md`.

Round 8 changed none of the seven Mermaid blocks (`extract_mermaid.py --check` read them identical to the sources of
`e3aedb25`) and none of the figures the case drawings read, so those nine differ from the drawings of `e3aedb25` only
in their titles' document identities, the PDFs' page size and, on the case plan, a footer that now wraps inside the
page and one label set on white. At `b7f96784` two Mermaid blocks differ from w3g's sources, the board interconnect's and the
power tree's dock edges (VIN_RAW on four 9 A pins at 14.10 A, EQ-16), and the case drawings read `c351115d`'s case
release (the plate's VHB lift 0.0, the as-coded plate and jacks moved; `case-drawings.md` names each input's commit).

## Findings the drawings surfaced

**At `b7f96784`** the build prints three disagreements (items 1, 3 and 4 below) and no netlist finding: item 2 is gone
because r8int4 re-declared the chain's pack for D-06, item 5 because W3B-R1 renamed board B's coin-cell net VBAT_RTC,
and item 6 because set 5 (board A stream w3a) made R74 and R133 the top legs of U16's and U19's enable dividers
(POE_UVLO, PD_UVLO), as the stage table's Enable column shows. Item 4 still prints because the SHORE_INPUT note names
the SMCJ33A as the clamp corrected away at `faf8c981` (stream w3de's rewording), which the check reads as a claim.

At `38dcd764`, reading the netlists against the declared energy chain (`power-tree.md`, first sections) finds the
same four disagreements with `v2/ecad/tools/pcb_energy_chain.yaml` as at `e3aedb25`, all in the chain file, none in a
circuit, plus one naming note:

1. Board P's chemical fuse F2 (Eaton SCF9550-30-05) is in series between FUSED and SCP_OUT; the chain has no F2 stage
   and runs its PACK_FETS stage from FUSED (PWR-F12; the re-declaration exists as a draft,
   `v2/docs/records/rv-pwr/pwr-chain-redeclaration.yaml`).
2. The chain's PACK_CELLS stage still reads "4S3P or 4S4P, about 200 Wh"; owner ruling D-06 made the pack one 4S3P block
   of Samsung 35E (about 145 Wh).
3. Stages B_PANEL_5V, B_HDMI_5V and B_QMX_5V take their prospective fault current from "board A's AP64500 buck U7"; board
   A's U7 is an LM5176PWPR making +5V_DEV, limited by its own current loop (ARCHITECTURE.md 4.1).
4. SHORE_INPUT's note names an SMCJ33A clamp; board E carries SMCJ40A and SMCJ40CA clamps since `faf8c981`.
5. Not a chain item: board B's net `VBAT` is its CR2032 backup, not board A's VBAT: one name on two boards, never joined.

They were handed to the owner of the energy chain as `v2/docs/records/hc4/energy-chain-disagreements.md`; nothing in the
chain file is changed here. The rebuild adds one netlist finding, printed by `power_tree.py` on every build:

6. **Board A's R74 (on POE_EN) and R133 (on PD_EN) each have both pins on one net.** They are the half of R4T-F3
   (`v2/docs/records/r4t/r4-decisions.md`) that round 8 did not close. Round 8 closed the other half on the PA and HF
   converters: R58 and R124 (10k 1%) now run from PA_EN and HF_EN to PA_UVLO and HF_UVLO over R59 and R125 (15k 1%)
   to GND, so U13 and U15 take 0.6 of their enable line. R74 and R133 do nothing, so the PoE and USB-C PD converters
   U16 and U19 sit on POE_EN and PD_EN directly, with R75 and R134 (10k 1%) as pull-downs: the way U5 (SLOT_EN2, R34
   100k to GND) and U7 (DEV_EN, R42 100k up to +3V3, S-08) are driven by design (`en_div=False` in `gen_sch_a.py`).
   U2 takes 0.68 of FE_RUN through its own supervisor network (R199 47k, R206 100k, C213 2.2n). `power-tree.md`
   prints how each LM5176's EN/UVLO pin is driven, read from the netlist on every build. For the board A author; no
   generator is changed here.
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

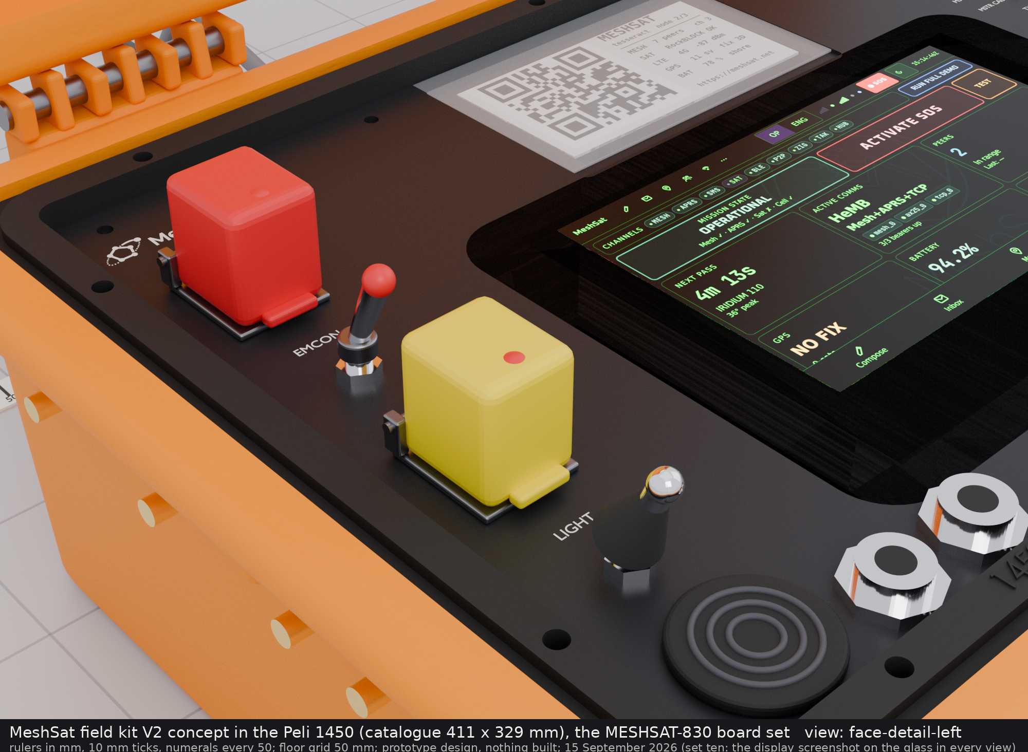
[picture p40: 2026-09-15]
v2/images/concept-1450/set-ten/08-face-detail-left.png

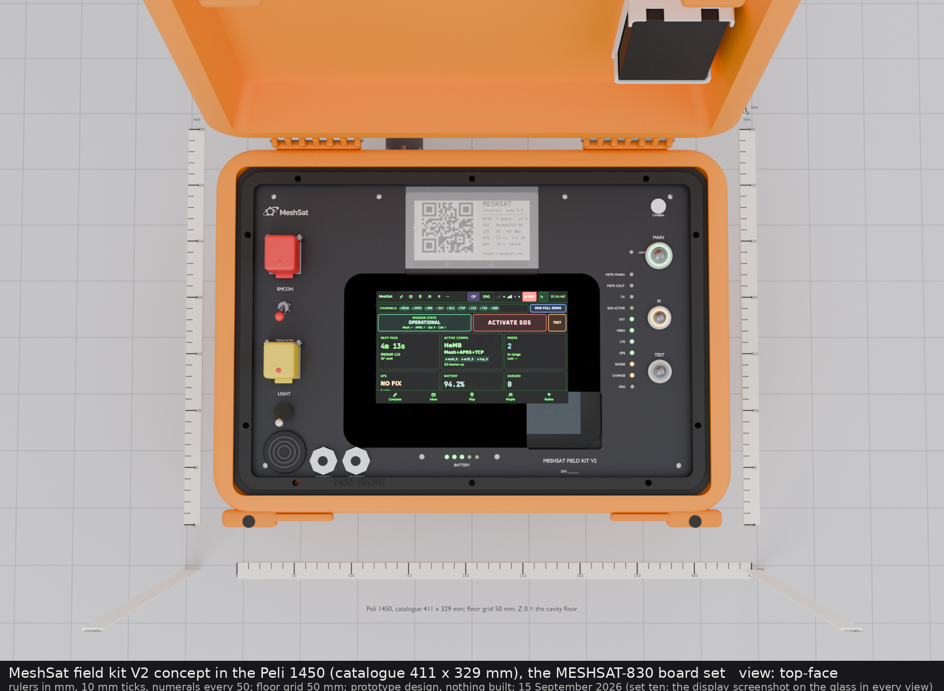
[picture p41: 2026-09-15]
v2/images/concept-1450/set-ten/07-top-face.png

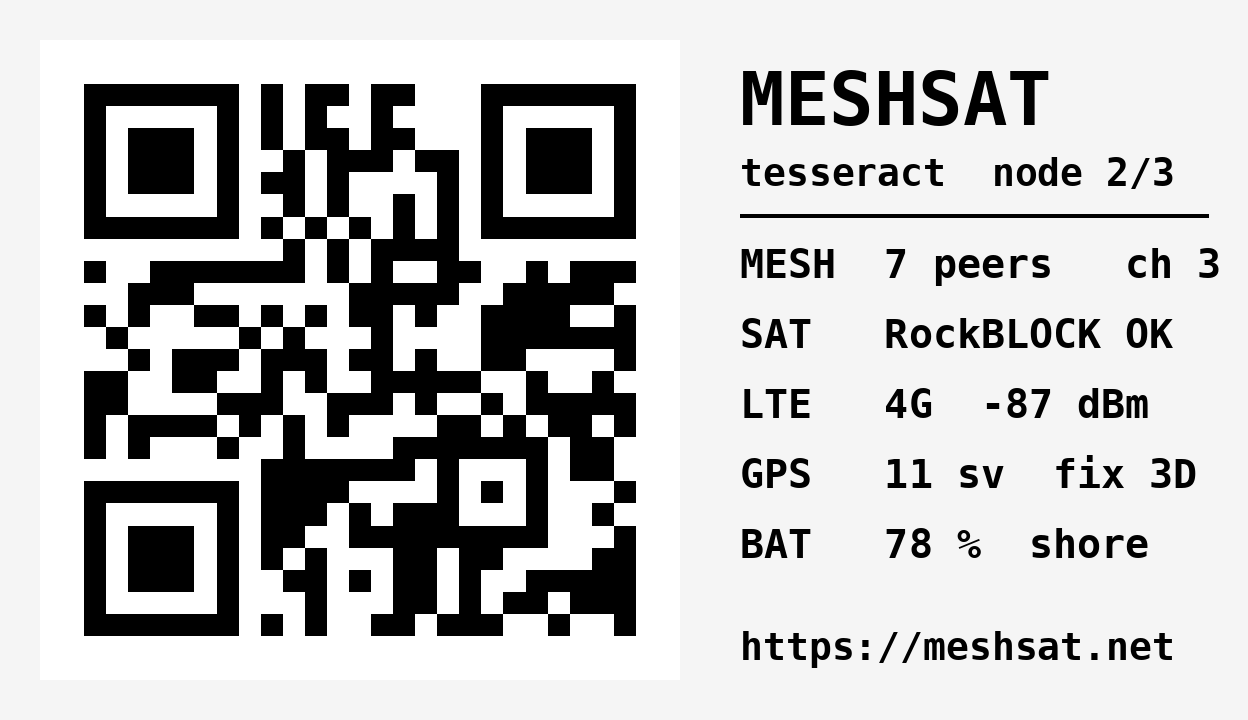
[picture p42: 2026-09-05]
v2/cad/render/epaper.png

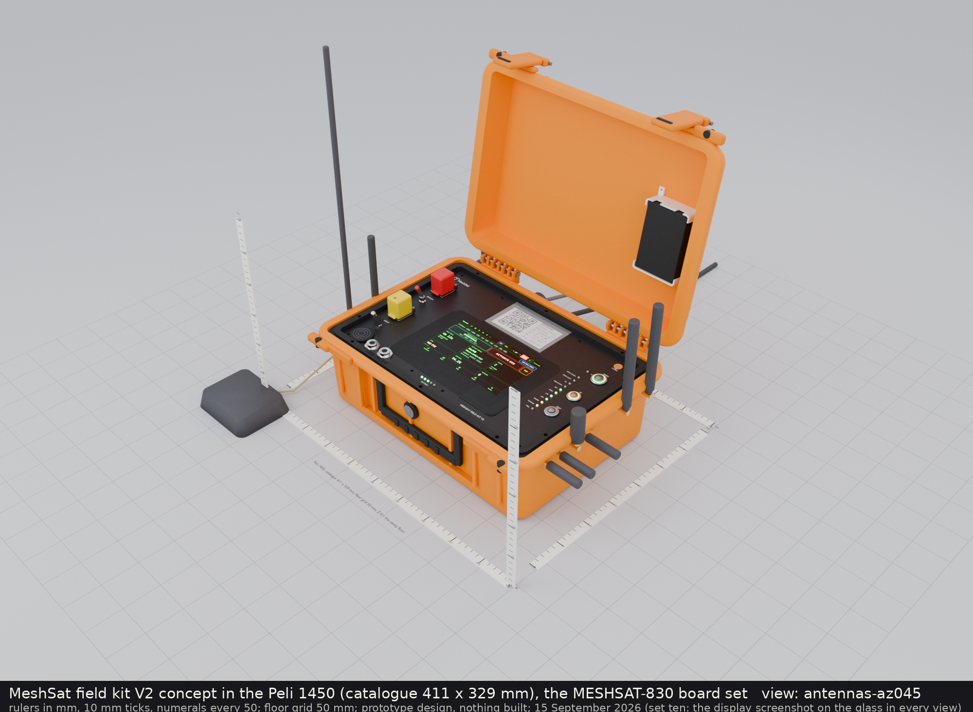
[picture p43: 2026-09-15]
v2/images/concept-1450/set-ten/18-antennas-az045.png

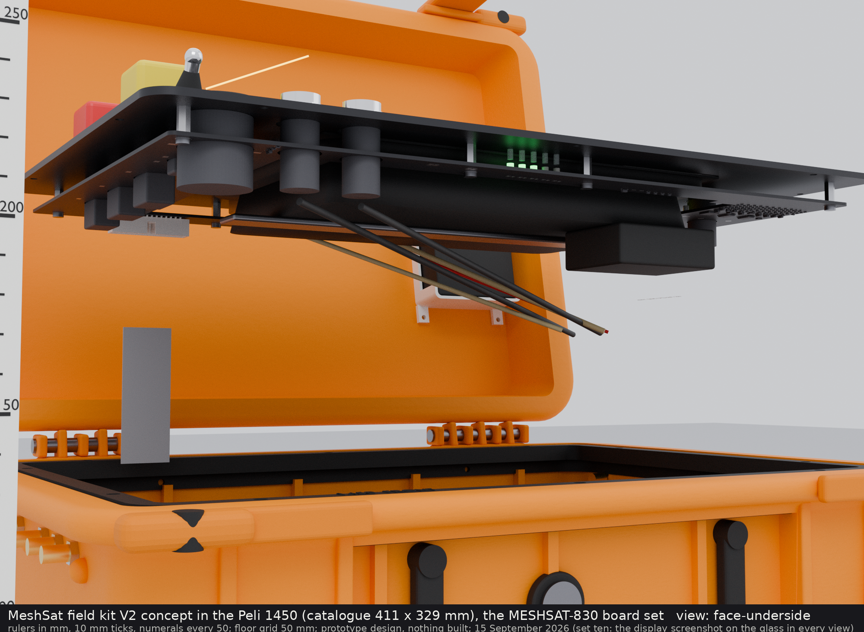
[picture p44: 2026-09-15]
v2/images/concept-1450/set-ten/10-face-underside.png

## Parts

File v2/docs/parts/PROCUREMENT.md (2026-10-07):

# Procurement constraints, supported alternatives and grade findings (pre-PCB layer 6)

Prototype design (MESHSAT-1357, closer hc6, 27 September 2026). Nothing has been built, bought for assembly, powered or
deployed. The order set stays quarantined (decision 41) and every purchase stays with the owner: this page orders
nothing, logs into nothing and puts nothing in a cart. Every stock figure is a reading of a public page at the time
given, and it is true only at that time.

**Judged at** main `53a98a71` (the six committed netlists, `v2/ecad/tools/lcsc_fill.py`, `v2/release/revA/order/JLC-CERTIFIED.tsv`):
round 8's boards A, D and E are integrated there; boards B, C and P are byte-identical to `e3aedb25`, where the layer 6
audit was taken. Quantities are per kit from the netlists, times five kits (the owner's "minimum 5 of each"). Board B's
round 8 part changes (the DS3231SN land, the U.FL codes, the key-B socket's locating holes) are in worktree `r8b`, not
on main; where one moves a row below it is said. Round 8's new codes on A and D (C2657885, C139409, C37593, C113780)
have no row in the certification table yet (the round 8 re-take left A32, D12 and E17 without a folder), so their
readings here are this page's own.

Companion pages: `v2/docs/parts/STM32H743-COMPATIBILITY.md` (the supervisor matrix), `v2/docs/parts/GRADE-CHECK.md`
(generated: every fitted active part and connector against the envelope, from `grade-sources.yaml` by
`grade_check.py`), and the readings in `v2/docs/parts/readings/`.

## 1. How the readings were taken

| Source | What was asked | When (UTC, 27 September 2026) | File |
|---|---|---|---|
| JLCPCB public parts API (the endpoint `jlc_certify.py:40` uses) | stock by LCSC code for 58 critical codes; keyword searches for alternatives | 00:02 to 00:20 | `readings/jlc-2026-09-27.json` |
| LCSC public product detail | model, stock, parameters, datasheet link for every code on a fitted BOM line (203 codes) | 00:04 to 00:07, 00:24 | `readings/lcsc-2026-09-27.json` |
| FindChips (Supplyframe's public aggregator page) | authorised and broker distributor offers for 51 order codes | 00:03 to 00:16 | `readings/findchips-2026-09-27.json` |
| Makers' pages and sheets | ranges, order codes and suffixes (Ground Control, Mill-Max, JST, Wurth, Pulse, Radiall, Preci-Dip) | 00:08 to 00:26 | filed in `v2/vendor/` (section 7) |
| JLCPCB public parts API, second reading | round 8's new codes on main and every constrained code of sections 2 and 3 again; keyword searches for HX6096NL | 03:59 to 04:06 | `readings/jlc-r8-main-2026-09-27.json` |
| Makers' pages, second pass | Pulse's product finder (HX6096NL sheet); URL checks of held documents (AsiaRF, Raspberry Pi, Radiall, Glenair, Xenarc) | 03:56 to 04:05 | section 7 |

FindChips repeats one stock figure across a distributor's packaging rows (cut tape, reel, Digi-Reel); the largest
figure per distributor is quoted, never the sum. A broker offer (Win Source, Chip Stock, Chip 1 Exchange, Unikey,
Bristol) is listed for completeness and is **not** a supported source for this prototype (HC6-SC-12).

## 2. The five constraints the audit named

### 2.1 Board P F2, the chemical fuse Eaton SCF9550-30-05 (C3670061)

- **Readings.** JLCPCB 0 (00:18:42Z), LCSC 0 (00:05:28Z); DigiKey 907 cut tape (283-SCF9550-30-05CT-ND), Avnet 0
  (lead time 12 weeks, MOQ 3000), Sager 0 (FindChips 00:13:37Z). Need 5.
- **Single source.** Eaton only; the SCF9550 order code fixes the cell count and the trip element, so no other code
  of the family is a drop-in: SCF9550-45-07 (C3667292, JLCPCB stock 10) is a 45 A part for a different cell count
  and stays a mismatch.
- **Alternatives, each a mismatch until the owed battery review R-BAT accepts it:** the Littelfuse ITV9550
  30 A family (`v2/vendor/battery/littelfuse-itv9550-30a.pdf`, SOURCES `pack-chemical-fuse-alternative`, evaluated
  and not fitted; every ITV9550 code at JLCPCB read 0 at 00:02:44Z), and the Dexerials SFK series
  (`v2/vendor/battery/dexerials-sfk-series-datasheet.pdf`, refused in round 4 for want of a published temperature range
  and land: `v2/vendor/vendor-status.txt`, FUSE-INTERPRETATION.md).
- **Grade.** "Operating temperature: -20 C to +60 C" (AT_LIMIT at the envelope's floor) and "Storage temperature:
  -10 C to +40 C < 90% RH, Storage duration: 1 year" (`v2/vendor/battery/eaton-scf9550-elx1135.pdf`, General
  specifications). The storage line reads like a shelf condition for the unmounted part; if it applies to the mounted
  fuse, it is narrower than the envelope's storage (-20 to +45 C) and the -33 C and +71 C margins. **Question for
  R-BAT and for Eaton (VENDOR_CONFIRMATION):** does the storage figure bind the assembled pack?
- **HC6-SC-9.** Buy SCF9550-30-05 from an authorised distributor and fit it as a hand-fit (consigned) line on board P,
  declared in board P's own `lcsc-allow.txt` (lcsc_fill reads only the board's own list, SOURCES
  `wrong_model_that_stands`); no alternative is adopted. Reverse if JLCPCB restocks before the order.

### 2.2 Board P U2, the second-level protector TI BQ7720700DSSR (C3681715)

- **Readings.** JLCPCB 3 (00:18:41Z), LCSC 3 (00:05:28Z): short of 5. DigiKey 2648 (cut tape, reel and Digi-Reel,
  FindChips 00:13:40Z). A search for the 250-piece reel BQ7720700DSST returned only DSSR offers.
- **Single source.** TI only; the "00" variant is the threshold set (OV 4.325 V, UV 2.25 V, OT 70 C) the pack design
  rests on; another BQ77207xx variant is a different protector, not an alternative.
- **Grade.** TA -40 to +85 C (`v2/vendor/battery/ti-bq77207.pdf`, Recommended Operating Conditions): INSIDE.
- **HC6-SC-9 (same rule).** Consign from an authorised distributor (DigiKey holds 2648) if JLCPCB still reads below 5
  at order time; the part does not change.

### 2.3 Board B Y1 to Y4, the 25 MHz crystal Yajingxin TAXM25M4RFBCCT2T (C164047)

- **Readings.** JLCPCB 3 (00:18:28Z, and again 3 at 04:00:03Z), LCSC 0 (00:04:46Z) against a need of 20 (four per kit: Y1 on the KSZ9897R, Y2 to
  Y4 on the three supervisors). FindChips shows LCSC with 19,150 at 00:13:45Z; LCSC's own API read 0 nine minutes
  earlier, so the aggregator's figure is taken as stale.
- **The criteria a replacement must meet.** The KSZ9897R's Table 6-12 (ESR at most 50 Ohm, +-50 ppm, 100 uW;
  `v2/vendor/cluster/ksz9897.pdf`, DS00002330E p.181) and the STM32H743's HSE criterion (gm_crit at or below
  Gmcritmax 1.5 mA/V, DS12110 Rev 11 Table 131). `STM32H743-COMPATIBILITY.md` section 7 computes both.
- **HC6-SC-3.** C9006 YXC X322525MOB4SI: JLCPCB basic library, 165,557 (00:18:29Z); YXC sheet ESR 50 Ohm, C0 3 pF,
  CL 12 pF, gm_crit 1.11 mA/V, pads 1/3 crystal and 2/4 ground (the `Crystal_GND24` symbol). Alternate C91750 Seiko
  Epson X1E0000210139, 6,098 (00:18:30Z), ESR 40 Ohm. The same land and load capacitors; the code change is board B's
  author's (`gen_sch_b.py:1150` and Y1's line).

### 2.4 Board D U2, the NiceRF SA868 order code (NOT_PINNED)

- **What the makers' documents give.** The held sheet V1.3 (`v2/vendor/nicerf/nicerf-sa868-datasheet-v1.3.pdf`) lists
  UHF 400 to 480 MHz, VHF 134 to 174 MHz and a 350 band as variants of one module and no order code. NiceRF's product
  page (Internet Archive capture of 2026-09-22 of
  `https://www.nicerf.com/item/2w-embedded-walkie-talkie-module-sa868`, fetched 00:02Z) offers "SA868 2W Embedded walkie
  talkie moduleV1.4", a newer sheet than the one held; its file host did not resolve from this host, and nicerf.com
  answered HTTP 403 to every product page.
- **The catalogue trap.** JLCPCB lists **SA868-U** (C3001507, stock 1, UHF) and **SA868S** (C52140339, stock 0, a
  different model). Neither is the part: the kit's APRS channel is 144.800 MHz, in the VHF variant only, and the S
  model is a substitution under condition 1.
- **HC6-SC-10.** The order code is **SA868-V** (NiceRF's band suffix, as its SA868-U and SA818S-V catalogue entries
  show). This is INFERRED from the maker's naming, not read in a NiceRF ordering table, so it carries a
  VENDOR_CONFIRMATION at purchase (the owner's) and the V1.4 sheet is owed. Reverse if NiceRF names the VHF variant
  otherwise.

### 2.5 Board B J_M2C2, the Quectel RM520N-GL order code (NOT_PINNED)

- **What exists.** Distributors list RM520NGLAA-M20-SGASA, -ESIM, -ESIM15, -PC15, -FC23 and RM520NGLAP-M20-SGASA
  (FindChips 00:03:33Z). Avnet describes -SGASA as the "MMWAVE M.2 FORM" standard SKU, RoHS true, lead time 13 weeks;
  the -ESIM variants carry an embedded SIM and read RoHS false; -PC15, -FC23 and the AP variant are not decoded by any
  held Quectel document. Stock: DigiKey 0 (MOQ 100, tray), Avnet 0; brokers only otherwise.
- **HC6-SC-11.** The order code is **RM520NGLAA-M20-SGASA**: the standard global SKU, a physical SIM through the
  socket's UIM lines (board B carries nano-SIM holders), RoHS. INFERRED from distributors' descriptions; a Quectel
  ordering document is owed and a VENDOR_CONFIRMATION goes with the purchase (the owner's, bought as a card).
- **Not an alternative.** RM520N-EU (the held hardware design V1.1 covers it) has five antenna ports (Table 32) against
  the GL's four, so the antenna plan changes.
- **Grade.** Operating -30 to +75 C, extended -40 to +85 C with 3GPP deviations (hardware design V1.1): INSIDE.

## 3. Single-source critical parts

"Critical" is SOURCES.yaml's own criterion (safety, a mission function, or a contested identity). Need = per kit x 5.
"Authorised" is the largest franchised-distributor figure FindChips showed. Every part here comes from one maker;
the "Alternative" column names what is supported and its state under condition 1.

| Part (order code) | Board, refs | Need | JLCPCB (UTC 00:18-00:19) | Authorised distributors (FindChips) | Constraint | Alternative and its state |
|---|---|---|---|---|---|---|
| ST STM32H743VIT6 (C114409) | B U41, U51, U61 | 15 | 4265 | DigiKey 0, Farnell 0, TME 39, Schukat 176 | revision V ONLY (SESSION L9T5-D11, 7 October 2026: HC6-SC-1's revision V or X narrowed, revision X NOT ADMITTED; no stock figure here reads a lot's revision, so an order names revision V; no query sent); franchised stock thin | STM32H743VIT6TR C5271084 (894, same part on reel): MATCH; STM32H753VIT6 C730206 (0): the first-named part, not needed |
| Microchip KSZ9897RTXI (C638299) | B U1 | 5 | 205 | DigiKey 4969, Avnet 44 | none | none needed |
| Diodes PI7C9X2G404SLBFDEX (C500767) | B U101, U201, U301 | 15 | 2770 | DigiKey 70 | franchised stock thin | PI7C9X2G304SL (held sheet) is a 3-port part: not a drop-in |
| TI TUSB8041IRGCR (C544686) | B U102, U202, U302 | 15 | 3180 | DigiKey 1304 | none | none needed |
| TI TMUXHS4212IRKSR (C3656912) | B U109, U209, U309 | 15 | 3909 | DigiKey 0, TME 0 | JLCPCB is the only franchised-grade stock read; the I suffix is the -40 to +105 C part | TMUXHS4212 without I is 0 to +70 C: not an alternative |
| TI TPS23861PWR (C93245) | B U5 | 5 | 26 | DigiKey 8813 | none | none needed |
| Pulse H5007NL (C6384935) | B T1 | 5 | 306 | DigiKey 6838, Farnell 632 | **grade OUTSIDE (0 to 70 C), and no PoE rating on its sheet while it carries the 802.3at feed** | HX6096NL, section 4 (HC6-SC-6) |
| Microchip ATECC608B-SSHDA-T (C1518769) | B U8 | 5 | 2342 | Avnet 8000, DigiKey 534 | the part choice waits on Z-EXP-A/B (FB-ZER-1, the owner's purchase) | SLB 9673 TPM 2.0 fallback, no JLCPCB stock (ARCHITECTURE.md line 1043 at `53a98a71`) |
| ADI DS3231SN#T&R (C9866) | B U9 | 5 | 4686 | DigiKey 5933 | the land at `e3aedb25` is SOIC-8 for a 16-pin part (round 8 r8b draws SOIC-16W) | none needed once r8b merges |
| TI BQ4050RSMR (C157570) | P U1 | 5 | 15945 | DigiKey 5311 | none | none needed |
| Keystone 3568 mini blade holder (no code) | A F1; E F1, F2, F3; P F1 | 25 | not placed by JLCPCB (through-hole) | not read: FindChips answered unrelated parts for the bare number (00:15:35Z) | hand-fit; route `v2/ecad/tools/jlc-handfit.txt:66` (DigiKey), allow lines on E and P since round 8 | none; range TBD (no Keystone sheet held, GRADE-CHECK.md) |
| TI BQ7720700DSSR (C3681715) | P U2 | 5 | **3** | DigiKey 2648 | short at JLCPCB | section 2.2 |
| Eaton SCF9550-30-05 (C3670061) | P F2 | 5 | **0** | DigiKey 907 | short at JLCPCB | section 2.1 |
| TI BQ25731RSNR (C2871872) | A U3 | 5 | 1137 | DigiKey 0 | franchised 0 | none needed while JLCPCB holds stock |
| TI LM5176PWPR (C442493) | A (7 stages) | 35 | 12309 | DigiKey 332 | none | none needed |
| TI TPS25740ARGER (C544309) | A U18 | 5 | 2949 | DigiKey 0 | franchised 0 | TPS25740B (held sheet) is another variant: a mismatch until compared |
| TI TPS259631DDAR (C2155778) | A, B (6 per kit) | 30 | 4423 | DigiKey 2576 | none | none needed |
| ADI LTC2954ITS8-1#TRPBF (C2657885, round 8, on main) | A U1 | 5 | **0** (00:18:48Z and 03:59:54Z) | DigiKey 4807 | **short at JLCPCB**; the code the design had before, #TRMPBF (C580654, 197), is not in the maker's order table and stays a condition 1 mismatch (SOURCES `power-button-controller`, `update_r8a`) | consign #TRPBF from DigiKey (HC6-SC-9); the part does not change |
| TI SN74AUP1G08DBVR (C139409, round 8) | A U35 to U38, the PA and HF rails' EMCON gates | 20 | 12,485 (03:59:56Z) | not read | none | none needed; another maker's 74AUP1G08 would be a substitution under condition 1 |
| TI ADS1115IDGSR (C37593, round 8) | D U22, the PA flange temperature ADC | 5 | 33,574 (03:59:57Z) | not read | TI only | none needed |
| ADI LT8705AEUHF#TRPBF (C674164) | E U5 | 5 | **3** | DigiKey 2438 (reel), 155 (#PBF tube) | **short at JLCPCB** (not named by the audit; found here) | LT8705AEUHF#PBF is the same part in a tube (the ordering table of the sheet LCSC serves lists #PBF and #TRPBF on one row): MATCH; consign from DigiKey |
| Quectel LG290P03AAMD (C29781241) | B U11 | 5 | 73 | DigiKey 35 | thin | none needed at 5 kits |
| Ebyte E22-900M30S (C411294) | B U12 | 5 | 551 | none franchised | Ebyte only | none needed |
| Ebyte E72-2G4M20S1E (C5352930) | B U13, U14 | 10 | **0** | none | **short at JLCPCB** (not named by the audit; found here) | Ebyte direct as a hand-fit module; no other maker makes this pin-out |
| Amphenol 10164227-1004A1RLF (C7435219) | B (6 receptacles) | 30 | 1238 | DigiKey 66 | JLCPCB is the stock | none needed |
| TE 2199119-3 (C590866) | B J_M2C2 | 5 | 1427 | DigiKey 8926 | land holes owed on main (S-12, r8b draws them) | none needed |
| TE 2199230-4 (C2977809) | B J_M2C1, J_M2C3 | 10 | 6464 | Farnell 7656 | none | none needed |
| TI TCAN334DR (C2871143) | B (6) | 30 | 479 | DigiKey 0, Farnell 317 | none | TCAN334GDR (5 Mbps, same pins) is not needed at 1 Mbps |
| Radiall R222M00720 (no code) | A J_BM1 to J_BM11 | 55 | not in catalogue | DigiKey 1335 | hand-fit; Radiall only | none (the blind-mate pair is a Radiall system) |
| Radiall R222M80500 (dock cable plugs) | dock block, one per receptacle | 55 | not in catalogue | DigiKey 349 as R222M80500W, 0 as R222M80500 | Radiall only | R222M80500W: "Packaging ... Unit 'W' option" on Radiall's own TDS p.2, so MATCH (packing) |
| Preci-Dip 813-S1-012-10-016101 (no code) | A J_DOCK | 5 | not in catalogue | DigiKey 18 (JRH listing), 0 (Preci-Dip listing) | **Preci-Dip only, 18 units seen** | none adopted: another spring connector is a different height and stroke (a mismatch, and the dock gap rule of 32.18 rests on it) |
| Mill-Max 0858-0-15-20-82-14-11-0 (no code) | A J_CP1-4, J_CN1-4 | 40 | not in catalogue | DigiKey 18646, Farnell 1401 | hand-fit (HC6-SC-8) | none needed; J_PRE1's longer pin has no order code (NOT_PINNED) |
| Raspberry Pi CM5108064 | B, three per kit (bench) | 15 | not in catalogue | Farnell 0, TME 0 | owner-side purchase through Raspberry Pi resellers | CM5108064B listed by Farnell (0): suffix not decoded |
| Ground Control RockBLOCK 9704 SMA | B, bench | 5 | not in catalogue | none listed | maker only; the maker's page publishes no order code | none |
| Lime Microsystems LimeSDR Mini v2 (v2.4) | B bay, bench | 5 | not in catalogue | none listed | **grade OUTSIDE (0 to 70 C)** | section 4 |
| AsiaRF AW7915-AED | B, two per kit (bench) | 10 | not in catalogue | none listed | **grade OUTSIDE (0 or -10 to 70 C)** | section 4 |
| NiceRF SA868-V | D U2 (bench) | 5 | SA868-U only (wrong band) | none | section 2.4 | none |
| Quectel RM520NGLAA-M20-SGASA | B J_M2C2 (bench) | 5 | not in catalogue | DigiKey 0, Avnet 0 | section 2.5 | none |
| Xenarc 709GNK | face plate | 5 | not in catalogue | DigiKey 6 | thin | none |
| Mitsubishi RA30H1317M1 | face plate | 5 | not in catalogue | brokers only | Mitsubishi only; the -501 and -101 suffixes the brokers list are not decoded | none; a qualified RF review should name the suffix |
| Amphenol PolyPhaser GTH-SFF-AL | wall | per jack | not in catalogue | Pasternack 0 | maker only | none |
| Glenair 233-370 USB feed-through | wall | 5 | not in catalogue | FindChips returned unrelated parts | made to order by Glenair | none |

## 4. Grade findings that need a decision (from `GRADE-CHECK.md`)

`GRADE-CHECK.md` judges 146 identities on the boards at `53a98a71` (every coded active part and connector by its code, and every
uncoded line by footprint; three of them are copper with no component) and 19 modules, cells and wall parts. Its findings:

| Finding | Part | Evidence | What it holds | Session recommendation |
|---|---|---|---|---|
| OUTSIDE, cold; PoE rating absent | Pulse H5007NL, board B T1 | "Operating Temperature 0 C to 70 C" (`v2/vendor/pulse/pulse-h5007nl.pdf` p.1). T1's media-side centre taps carry the 802.3at feed (`POE_P` on pin 24, `POE_DRAIN` on pin 21; `gen_sch_b.py:866-869`), and the HC500.O sheet states no DC current or voltage rating for any part it lists; Microchip's Table 7-2 lists H5007NL for data only | the wall Ethernet port below 0 C, and the PoE out function at any temperature (condition 1: a part not documented for a function the design gives it is a mismatch until proven) | **HC6-SC-6: HX6096NL** (Pulse; C5339289 HX6096NL, JLCPCB 146, or the reel HX6096NLT C5359044, 323, both at 04:05:50Z). Its sheet (`v2/vendor/pulse/pulse-hx6096nl-datasheet-rev-a.pdf`, filed tonight) reads "OPERATING TEMPERATURE -40 C - +85 C", "DC CURRENT/VOLTAGE RATING 720 mA, @ 57 V (CONTINUOUS)" and "MEETS IEEE 802.3 SPECIFICATION"; its pin numbering is T1's own (chip side TCT1 1 ... TD4 11/12, media side MCT1 24 ... MX4 14/13) and its suggested land (24 x 0.76 mm on 1.27 mm, rows 12.70 mm inner and 16.51 mm outer) is the one `meshsat:Pulse_H5007NL` already draws, so no pad moves. The body grows from 17.53 x 12.20 x 5.51 to 18.16 x 12.2 x 6.60 mm (placement and stack-height input). Residual for R-PWR (the PoE PSE): Microchip's Table 7-1 asks 350 uH minimum at 8 mA; Pulse guarantees 350 uH at +25 C with 24 mA of bias and 300 uH across -40 to +85 C. The generator line (`gen_sch_b.py:869`) is board B's author's. **Withdrawn:** HX5008NL, which this page first recommended from Microchip's Table 7-2, has no PoE rating in HC500.O and needs a new land; HX5004NL has neither a PoE rating nor an OCL figure. The CND-tek HX6096NLTP-CND (C47575006) is another maker's part and is not the recommendation (HC6-SC-12) |
| OUTSIDE, cold and storage | LimeSDR Mini v2, v2.4 | "Operating Temperature 0 C to +70 C, Commercial-grade; Storage Temperature 0 C to +70 C" (`v2/vendor/limesdr/myriadrf-limesdr-mini-2-0-page-20260925.html`) | the SDR receiver below 0 C, and its storage in the kit below 0 C | open: (a) an industrial-grade USB SDR in the same bay (a part search and the bay's L7 fit are owed), (b) a carve-out in OPERATING-ENVELOPE.md, which narrows the kit and is not the session's to take, (c) warming the bay before use, which needs a heat source the design does not have. The SDR is not in D-01's core (CONOPS 2a), so this holds no core acceptance; it does hold NEED-07 for that function |
| OUTSIDE, cold | AsiaRF AW7915-AED (two) | "Temperature Operating: 0 C ~ +70 C" (`v2/vendor/wifi/asiarf-AW7915-AED_V1.pdf`); the maker's page of 26 September reads -10 C ~ +70 C | the kit-to-kit WiFi link below 0 C (or -10 C); CONOPS 2a exercises it through IOHA test A11 | open: an extended-temperature M.2 2230 E-key card with the mt76 driver the P2P mission needs (a search is owed; the socket and land do not change, so the choice can wait until before purchase without touching layout); the carve-out option is not the session's |
| AT_LIMIT, cold (no margin at -20 C) | CM5 module, Xenarc 709GNK, Wurth 692122030100 USB 3 A, SGP41 (also +55 C against 51 C of air), C&K ATP16 and ATP19 switches, Floyd Bell sounder class, SCF9550, GCT SIM8060 (one of its two sheets), Amass XT60-M, Bulgin PX0833 | `GRADE-CHECK.md` | nothing at the envelope; the -33 C qualification margin is a survive-and-recover line | none: the envelope is met; each is reported for the margin tests of TEST-PLAN E3/E4 |
| TBD, no range read | Keystone 3568 and 3034 holders, the sixteen 3 mm panel LEDs, the headset jacks, the J_PRE1 pin, commodity pin headers, the Molex 208658 HDMI receptacle (molex.com and LCSC's copy did not answer), SS14 (C51897884, no sheet), QMX, the fans, the pack cells, the CR2032 cell, the sensor modules on headers | `GRADE-CHECK.md` | NEED-07 for each; none is a mission part except the pack cells (owed by the pack pick) | the NOT_PINNED ones get a range when they get an order code |

## 5. Interface parts identified tonight (session picks)

| Id | Pick | Why | Reversal |
|---|---|---|---|
| HC6-SC-7 | IDC box headers: Wurth WR-BHD 61202621621 (2x13, JLCPCB C17586777), 61201621621 (2x8, C5364137), 61201021621 (2x5, C4355000), all -40 to +105 C, 3 A per contact; mating IDC sockets WR-BHD 61202623021, 61201623021, 61201023021 (1 A per contact, -40 to +105 C); flat cable WR-CAB 63912615521CAB, 63911615521CAB, 63911015521CAB (1.27 mm, 28 AWG, 1 A, -25 to +105 C, UL AWM 2651 105 C 300 V). Board C's SMD 2x13 header: XFCN BH254VS-26P (C48687640, LCSC parametric -40 to +105 C) | one maker for header, socket and cable, with sheets fetched from we-online.com (section 7); the ribbon's 1 A per conductor is the figure the interface capacity rows (layer 5) must be checked against | a different maker if the land comparison (below) fails; the SMD header is the weakest pick (no maker sheet read) |
| HC6-SC-8 | Mill-Max 0858-0-15-20-82-14-11-0 for J_CP1-4 and J_CN1-4 (82 spring, "12 Amp High Force" on Mill-Max's page; the 085X family is "Continuous 9 amps @ 10 C temperature rise", catalogue page 28) | the part the land was drawn for (`respin-footprints-2026-09-04.md` section 5), DigiKey 18,646 | none planned |
| HC6-SC-12 | buy only from JLCPCB/LCSC stock or franchised distributors; no broker stock | counterfeit and relabelled-revision risk, which F1 (silicon revision) makes concrete for the supervisors | none |

**Land comparisons these picks create (CMP-002's identity-and-land half, owed at layout entry):** the Wurth
WR-BHD recommended hole pattern against KiCad's `IDC-Header_2x13_P2.54mm_Vertical_NarrowPad` (and the 2x5, 2x8
lands); the XFCN drawing against `IDC-Header_2x13_P2.54mm_Vertical_SMD`; the Mill-Max 0858's ".044 in (1,118 mm)"
mounting hole for its ".040 in (1,016 mm)" tail against the land's 1.3 mm drill (`respin-footprints-2026-09-04.md`
section 5 took its hole from the strip page's 1.32 mm): a solder mount tolerates the larger hole, but the pin's
squareness then rests on the assembly fixture, which ASSEMBLY.md should say.

## 6. Session choices on this page

HC6-SC-3 (crystal), HC6-SC-6 (magnetics), HC6-SC-7 (IDC), HC6-SC-8 (Mill-Max), HC6-SC-9 (consign SCF9550 and
BQ7720700), HC6-SC-10 (SA868-V), HC6-SC-11 (RM520NGLAA-M20-SGASA) and HC6-SC-12 (sources) are the session's, taken
under the owner's standing rule of 26 September 2026 because each follows from the makers' documents and no owner
judgement is standing; each names its reversal above. HC6-SC-1, -2, -4 and -5 are on `STM32H743-COMPATIBILITY.md`.
None changes a requirement, a function or a protection; the generator lines that would carry HC6-SC-3, -6, -7 and -8
belong to the board authors and are listed in `drafts/hc6/README.md` of the worktree that wrote this page.

## 7. Documents filed tonight

| File | What | sha256/16 | Source |
|---|---|---|---|
| `v2/vendor/st/st-stm32h743xi-datasheet-rev11.pdf` | ST DS12110 Rev 11 (13 January 2026) | `f6e620179006c8c4` | Internet Archive, capture 20260827112637 (gzip body decompressed); capture 20260318060051 identical |
| `v2/vendor/st/st-rm0433-rev8.pdf` | ST RM0433 Rev 8 (January 2023), 40.7 MB | `9ba54135736a47a3` | Internet Archive, capture 20251014013150 |
| `v2/vendor/st/st-es0392-rev15.pdf` | ST ES0392 Rev 15 (September 2025) | `effe23b2b79ec4ee` | Internet Archive, capture 20260526205148 (gzip body decompressed) |
| `v2/vendor/connectors/jst-vh-catalogue.pdf` | JST VH connector catalogue (PDF of 9 January 2026) | `d51e669c597988b2` | https://www.jst-mfg.com/product/pdf/eng/eVH.pdf, 00:21Z |
| `v2/vendor/connectors/wurth-wr-bhd-box-header-61202621621.pdf`, `-61201621621.pdf`, `-61201021621.pdf` | Wurth WR-BHD box headers (dated 2026-08-30) | `38509e478ba394d0`, `0df87add7e40d43c`, `dbaa4765e57457ac` | https://www.we-online.com/components/products/datasheet/<code>.pdf, 00:20Z |
| `v2/vendor/connectors/wurth-wr-bhd-idc-socket-61202623021.pdf`, `-61201623021.pdf`, `-61201023021.pdf` | Wurth WR-BHD female IDC connectors (dated 2022-08-30) | `6f7254b5bcf6f837`, `9477ffdc02af6355`, `259dc513fa09e911` | as above |
| `v2/vendor/connectors/wurth-wr-cab-ribbon-63912615521cab.pdf`, `-63911615521cab.pdf`, `-63911015521cab.pdf` | Wurth WR-CAB flat cable (dated 2026-08-21) | `fdee657377aed9ac`, `b076f824f67b9ee7`, `4b4b78e0c17b7f1d` | as above |
| `v2/vendor/connectors/wurth-wr-com-usb3-a-692122030100.pdf` | Wurth 692122030100 USB 3.0 A (board B J_LIME's land) | `df28a01bf0fb46ac` | as above |
| `v2/vendor/connectors/millmax-0858-product-page-20260927.html` | Mill-Max 0858 product page | `7a11ec390b01e69f` | https://www.mill-max.com/products/discrete-spring-loaded-pins/spring-loaded-pin-with-standard-tail/0858, 00:12Z |
| `v2/vendor/connectors/millmax-rugged-power-spring-pins-page28.pdf` | Mill-Max "Rugged, High Current Spring Pins" (catalogue page 28, 2014) | `8ef40cd98d95c653` | https://www.mill-max.com/sites/default/files/external/assets/2017-12/Rugged%20Spring%20Pins.pdf, 00:13Z |
| `v2/vendor/rockblock/groundcontrol-rockblock-9704-product-page-20260927.html` | Ground Control product page | `3ee56a034ace33a7` | https://www.groundcontrol.com/product/rockblock-9704/, 00:08Z |
| `v2/vendor/rockblock/groundcontrol-docs-rockblock-9704-specification-20260927.html` | Ground Control specification page | `30bad6e0074bea49` | https://docs.groundcontrol.com/iot/rockblock-9704/specification, 00:08Z |
| `v2/vendor/crystals/yajingxin-taxm25m4rfbcct2t-spec-2026-08-26.pdf` | Yajingxin specification of the fitted 25 MHz crystal | `cf02a0872e39ea73` | LCSC's datasheet link for C164047, 00:04Z |
| `v2/vendor/crystals/yxc-ysx321sl-x322525mob4si.pdf` | YXC YSX321SL (X322525MOB4SI) | `7bc18549e407d8e3` | LCSC's datasheet link for C9006, 00:05Z |
| `v2/vendor/crystals/epson-tsx-3225-x1e0000210139.pdf` | Seiko Epson FA-238/TSX-3225 sheet | `4e9c0baa33e30d2d` | LCSC's datasheet link for C91750, 00:05Z |
| `v2/vendor/pulse/pulse-hx6096nl-datasheet-rev-a.pdf` | Pulse HX6096NL, datasheet rev. A (07/30/15), 3 sheets, raster | `76b47ba60ec87752` | https://productfinder.pulseeng.com/doc_type/WEB301/doc_num/HX6096NL/doc_part/HX6096NL.pdf, 04:05:06Z (declared in `vendor-noindex.txt`) |

The held RockBLOCK 9704 data sheet (`v2/vendor/rockblock/rb9704-datasheet-RB9704-001-JUN26.pdf`) was re-fetched from
https://www.groundcontrol.com/wp-content/uploads/2026/07/RockBLOCK-9704-Data-Sheet.pdf at 00:26Z and is byte-identical
(its currency is confirmed and its URL is now known). The Pulse sheet LCSC serves for HX5004NLT is byte-identical to the
held `pulse-h5007nl.pdf`. Three more held files came back byte-identical from their makers at 03:56Z to 03:57Z, which
records their URLs: `wifi/asiarf-AW7915-AED-datasheet.pdf` (AsiaRF's 260505 one-page sheet), `cm5/cm5-datasheet.pdf`
(datasheets.raspberrypi.com), `rf/radiall-smp-max-series-R222M-D1C004XEe.pdf` (radiall.com). Not confirmed: the Radiall
per-part data sheets and the Glenair sheets (both makers answered HTTP 403) and the Xenarc manual and drawing (served
through a script); the Internet Archive was offline at 03:57Z, so their currency stays unconfirmed. The sources.txt and vendor-status.txt lines for these files are drafts
(`drafts/hc6/vendor-lines.patch`), because both files are shared.
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

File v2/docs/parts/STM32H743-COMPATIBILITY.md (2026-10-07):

# STM32H743 compatibility matrix: board B's three I/O supervisors

Prototype design (MESHSAT-1357, pre-PCB layer 6, closer hc6, 27 September 2026). Nothing on this page has been built,
bought for assembly, powered or measured. It is a desk comparison of ST's own documents against the committed
schematic, made by the session; it is not a qualified engineer's review and not a test.

**The question (owner condition 1, CON-017, S-41, D-13).** The design first named the STM32H753VI for the supervisors
U41, U51 and U61 (`v2/docs/research-io-supervisor-2026-09-09.md:3-4`); the purchase code C114409 buys the
STM32H743VIT6, and owner ruling D-13 of 26 September 2026 accepted the H743 with software-verified boot as the
prototype's floor. Since `458b2873` the symbol, value and order line name the STM32H743VIT6
(`v2/ecad/tools/gen_sch_b.py:1145-1146`). Condition 1 says a substitution is a mismatch until it is shown compatible. This page is the
proof CON-017 clause (3) asks for: every pin, peripheral and electrical feature the schematic uses, read in the H743's
own documents, set against the H753 the design first named, and every H753-only unit checked for a dependence.

**Judged at** main `e3aedb25`: `v2/ecad/tools/gen_sch_b.py` sha256/16 `dedaf34ce285e5ff` (lines 281-289 the pin table,
1085-1158 the control plane) and the committed netlist `v2/ecad/pcb-b-compute-b19/out/pcb-b-compute.net` sha256/16
`669d02d07aeaae4b` (U41, U51 and U61 read pin by pin). The round 8 board B candidate in worktree `r8b` changes one net
on these parts (pin 33, PC5, reads `EMCON_SUP`, a 74LVC1G34 copy of `EMCON_HW`, EMCON finding L1); every pin number,
pin function and alternate function below is the same in that candidate (netlist compared pin by pin for all three
supervisors on 27 September 2026). Re-checked at main `53a98a71`, where round 8's boards A, D and E are integrated:
`gen_sch_b.py` and board B's netlist are byte-identical there (sha256/16 `dedaf34ce285e5ff` and `669d02d07aeaae4b`), so
every row below stands.

## 0. Verdict

| Clause | State | Evidence |
|---|---|---|
| CON-017 (1) the schematic, symbol and BOM name the STM32H743VIT6, pin map unchanged | MET (held since `458b2873`) | `gen_sch_b.py:1146`; netlist value of U41, U51, U61; `v2/docs/records/r4b/pin_parity.py` (100 of 100 pins agree between DS12110 Figure 5 and DS12117 Figure 4) |
| CON-017 (2) regeneration parity traced | MET (CON-017 evidence, clamp-symbol merge) | `v2/ecad/tools/pcb_requirements.yaml` CON-017 evidence |
| CON-017 (3) compatibility matrix of every peripheral and feature used, with DS12110 sources | **MET by this page** (sections 2 to 6) | DS12110 Rev 10 and Rev 11, RM0433 Rev 8, ES0392 Rev 15, AN4938 Rev 7 |
| CON-017 (4) the supervisor firmware builds for the STM32H743 | **OPEN, allocated to the firmware stage** (section 8): no supervisor firmware exists, and nothing the layout decides depends on it | none; proposed registry change in `drafts/hc6/apply_registry.py` |
| Dependence on an H753-only unit (CRYP, HASH, secure access mode, RSS, secure-only flash) | **NONE** in any requirement, generator line or feasibility page (section 5) | RM0433 Rev 8 Table 2, p.103 |

Seven findings the design must carry. None changes a pin, a land or a net; they are procurement, firmware and
record obligations, each placed at the stage where its evidence can exist:

- **F1, silicon revision (procurement and firmware).** The design uses both FDCAN controllers. ES0392 Rev 15 section
  2.24.2 ("Wrong data may be read from message RAM by the CPU when using two FDCANs", workaround: none) is present on
  silicon revision Y and W and absent on X and V; so are 2.2.8 (PCROP areas may be unprotected, which touches D-13's
  verified boot) and 2.2.14 (leakage when an input is above VDD, which is the dark-controller case of IOHA A4). The
  supervisors must be revision V or X: marking V or X, REV_ID 0x2003 or 0x2001 in DBGMCU_IDC (ES0392 Table 2, p.1;
  RM0433 p.3208) [the erratum's bound; the selection inside it is revision V ONLY, marking V and REV_ID 0x2003, SESSION L9T5-D11 of 7 October 2026 (record l9t5, `T10-ROUND5.md` section W133): revision X is NOT ADMITTED and a lot marked X is refused]. Checked at goods-in (ASSEMBLY) and read by the firmware at boot. Session choice HC6-SC-1, narrowed to revision V by SESSION L9T5-D11.
- **F2, the kit bus (firmware contract).** A supervisor is an I2C target on the same SDA and SCL as the expanders, the
  PoE controller, the holdover clock and the secure element (`ARCHITECTURE.md` 5.5). ES0392 2.19.9 ("Transmission
  stalled after first byte transfer", a state in which the peripheral is stalled in target mode with clock stretching
  enabled) would hold SCL and stop the whole bus; 2.19.3 needs the I2C kernel clock at 10 MHz or more in Fast mode;
  2.19.10 holds SDA low if SMBus timeouts are used in target mode. Obligations in section 6. Session choice HC6-SC-2.
- **F3, the HSE crystal (part choice).** The fitted 25 MHz C164047 meets the oscillator criterion on its maker's own
  sheet (gm_crit 0.67 mA/V against Gmcritmax 1.5 mA/V), but it is NO_STOCK (3 against 20) and LCSC's parametric for it
  states 80 Ohm where the maker's sheet states 30 Ohm maximum. Any replacement is chosen by the same computation;
  section 7 gives it for two stocked candidates. Session choice HC6-SC-3 (recommendation to board B's author).
- **F4, document currency.** DS12110 Rev 10 (March 2023), the revision every record cites, is superseded by Rev 11
  (13 January 2026), which updated the pin table, the alternate function table, the operating conditions, VCAP, the
  I/O static characteristics and the I2C characteristics. Every row used here was re-read in Rev 11: no used pin,
  alternate function or relied-on value changed (sections 2 and 3). Rev 11 is filed.
- **F5, rev Y tables cited for a rev V part.** DS12110 carries two electrical sections, section 6 for silicon revision
  Y and section 7 for revision V. `gen_sch_b.py:1020` and `:1108-1114` cite Rev 10 Tables 21, 22, 24 and 60, which are
  the revision Y section. The revision V tables (Rev 10 Tables 119, 120, 122, 157; Rev 11 Tables 109, 110, 112, 147)
  give the same figures the design relies on: TT_xx input 4.0 V absolute maximum, "Positive injection is not possible
  on these I/Os", and TT_xx leakage +-250 nA (section 4). No circuit change; the citation should name section 7 (a
  comment for board B's author, recorded in `drafts/hc6/README.md`).
- **F6, the watchdog starts in hardware (provisioning).** `ARCHITECTURE.md` 6.1 has "option-byte start TBD (RM0433 not
  held)". RM0433 is now held: IWDG1_SW = 0 in the user option bytes makes "the watchdog ... automatically enabled at
  power-on" (RM0433 Rev 8 p.179; FLASH_OPTSR bit 4, p.214), clocked by the LSI and "active even if the main clock
  fails" (p.1894). Session choice HC6-SC-4: hardware watchdog, IWDG frozen in neither Stop nor Standby, written at
  provisioning with the other option bytes.
- **F7, the records disagree.** `v2/vendor/SOURCES.yaml` (io-supervisor-mcu, `update_45bde541`: identity MATCH, reopen
  conditions settled), `ARCHITECTURE.md:586` at `53a98a71` ("Owner condition 1 is not closed by the text"), `ARCH-PCB-B-IOHA.md`
  section 6 ("baseline 3x STM32H753", I2C on PB1/PB2 as an open finding) and section 10a (the rename "has not been
  done yet"), and S-41 (supervisor addresses 0x30 to 0x32, where `ARCHITECTURE.md` 5.5 took 0x34 to 0x36 under
  I3-F01) describe four different states. Patches that make them agree with this page are in `drafts/hc6/`.

## 1. Documents read

| Document | Revision | File in this tree | sha256/16 | Source and currency |
|---|---|---|---|---|
| ST DS12110, STM32H742xI/G STM32H743xI/G datasheet | Rev 10, 30 March 2023 | `v2/vendor/st/st-stm32h743xi-datasheet.pdf` | `9b27d1d993a8bc5b` | Wayback copy (st.com refuses this host); **superseded by Rev 11** |
| ST DS12110 | **Rev 11, 13 January 2026** (PDF dated 15 to 21 January 2026) | `v2/vendor/st/st-stm32h743xi-datasheet-rev11.pdf` (filed now) | `f6e620179006c8c4` | `https://web.archive.org/web/20260827112637id_/https://www.st.com/resource/en/datasheet/stm32h743vi.pdf`, fetched 2026-09-26T23:51Z; the archive served it gzip-encoded and the filed file is the decompressed body; the capture of 2026-03-18 (`20260318060051id_`) is byte-identical; st.com answered this host with an HTTP/2 INTERNAL_ERROR at 2026-09-26T23:49Z |
| ST DS12117, STM32H753xI datasheet | Rev 9, March 2023 | `v2/vendor/st/st-stm32h753xi-datasheet.pdf` | `3bf346d8a511843a` | Wayback copy; the newest archived capture is of 2023-06-08, so a newer revision is not excluded (the H753 is not fitted; it is read only for what it adds) |
| ST RM0433, STM32H742, STM32H743/753 and STM32H750 reference manual | **Rev 8, January 2023** (3353 pages) | `v2/vendor/st/st-rm0433-rev8.pdf` (filed now, 40.7 MB) | `9ba54135736a47a3` | `https://web.archive.org/web/20251014013150id_/https://www.st.com/resource/en/reference_manual/rm0433-stm32h742-stm32h743753-and-stm32h750-value-line-advanced-armbase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`, fetched 2026-09-26T23:50Z; newest capture 2025-10-14, still Rev 8 |
| ST ES0392, device errata | **Rev 15, September 2025** | `v2/vendor/st/st-es0392-rev15.pdf` (filed now) | `effe23b2b79ec4ee` | `https://web.archive.org/web/20260526205148id_/https://www.st.com/resource/en/errata_sheet/es0392-stm32h742xig-stm32h743xig-and-stm32h753xi-device-errata-stmicroelect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`, fetched 2026-09-26T23:52Z, served gzip-encoded, filed decompressed |
| ST AN4938, hardware development | Rev 7, 29 October 2024 | `v2/vendor/st/st-an4938-rev7.pdf` | `217b5dcbfdd27cec` | Wayback copy of 2025-07-26 (SOURCES.yaml io-supervisor-mcu) |

Rev 11 reads "refer to RM0399 reference manual" in its I2C section (p.297); RM0399 is the STM32H745/755/747/757 manual,
so that is a documentation slip, and RM0433 is the manual for this part (its own title and ES0392's applicability line).

## 2. Identity, package and grade

| Item | STM32H743VIT6 (fitted) | STM32H753VIT6 (first named) | Verdict |
|---|---|---|---|
| Ordering code | V = 100 pins, I = 2 MB flash, T = LQFP, 6 = -40 to +85 C (DS12110 Rev 11 section 9, p.346; Rev 10 p.348) | same scheme (DS12117 Rev 9 section 9) | the code buys the part the land and the pin table describe |
| Package | LQFP-100 14 x 14 mm, 0.5 mm pitch; pinout Figure 5, p.55 of both revisions | DS12117 Figure 4, p.55 | 100 of 100 pins agree (`records/r4b/pin_parity.py`, RECORDED) |
| Operating range | TA -40 to +85 C at maximum power dissipation, TJ -40 to +125 C (105 C at VOS0) (Rev 11 Table 112, p.210) | same | against `v2/ecad/tools/pcb_envelope.yaml`: -20 C floor and 51 C worst inside air (part_temps.py's bar): **INSIDE**, 34 K below the TA limit |
| Storage | TSTG -65 to +150 C (Rev 11 Table 111, p.208) | same | covers the -33 C and +71 C qualification margins |
| Stock | C114409 CERTIFIED (`JLC-CERTIFIED.tsv:582-584` at `53a98a71`, the reading of 26 September 2026: 4270); JLCPCB 4265 at 2026-09-27T04:00:07Z; tape-and-reel C5271084 | C730206 stock 0 | see `v2/docs/parts/PROCUREMENT.md` |

## 3. Every pin the schematic uses

Net names are supervisor A's (U41); B and C carry the same functions on their own `IOCB_`/`IOCC_` nets, the shared
`HB1..3`, `BSEL1..3`, `WIFI_SEC`, `EMCON_HW`, `SCL`, `SDA`, and their own `SEL`, `HUBRST` and `WSEC` bits. I/O
structure is DS12110 Table 9's column, read in Rev 10 and in Rev 11 (pp. 64 to 88): identical for every row. Pins
not listed are unconnected (56) or supplies (14).

| Pin | Name | I/O structure | Net (U41) | Use | Function and mode | Source (DS12110 Rev 11; Rev 10 in brackets) | Verdict |
|---|---|---|---|---|---|---|---|
| 12 | PH0 | FT | `IOCA_XI` | HSE crystal | OSC_IN, additional function | Table 9; section 7.3.7 Table 131 p.229 | MATCH (section 7 for the crystal) |
| 13 | PH1 | FT | `IOCA_XO` | HSE crystal | OSC_OUT | as above | MATCH |
| 14 | NRST | RST | `IOCA_RST_n` | reset, 10 k to 3V3, 100 nF to GND | bidirectional, internal pull-up RPU 30 to 50 k | Table 152 p.248 (Table 162) | MATCH; the 100 nF is Figure 74's "Recommended NRST pin protection" (0.1 uF, p.248), and the external 10 k sits in parallel with RPU |
| 22 | PA0 | FT_a | `SEL1_A` | voted bank 1 select, output | GPIO push-pull | Table 9 | MATCH |
| 23 | PA1 | FT_ha | `SEL2_A` | voted bank 2 select, output | GPIO | Table 9 | MATCH |
| 24 | PA2 | FT_a | `SEL3_A` | voted bank 3 select, output | GPIO | Table 9 | MATCH |
| 25 | PA3 | FT_ha | `HUBRST1_A` | voted hub 1 reset, output | GPIO | Table 9 | MATCH |
| 28 | PA4 | TT_a | `HUBRST2_A` | voted hub 2 reset, output | GPIO; injection 0/0 on PA4, PA5 (Table 110) | Table 9, Table 110 p.208 | MATCH as an output (100 k pull-down only; nothing drives it from outside) |
| 29 | PA5 | TT_ha | `HUBRST3_A` | voted hub 3 reset, output | GPIO; as PA4 | as PA4 | MATCH |
| 30 | PA6 | FT_a | `HB1` | module 1 heartbeat, input | GPIO input | Table 9 | MATCH |
| 31 | PA7 | TT_a | `HB2` | module 2 heartbeat, input | GPIO input, TT: 4.0 V absolute | Table 9, Table 109 | MATCH (section 4) |
| 32 | PC4 | TT_a | `HB3` | module 3 heartbeat, input | GPIO input, TT | as PA7 | MATCH |
| 33 | PC5 | TT_a | `EMCON_HW` (r8b: `EMCON_SUP`) | EMCON state, input only (round 6 O-06) | GPIO input, TT | as PA7 | MATCH; firmware keeps it an input (section 6) |
| 34 | PB0 | FT_a | `IOCA_LED_A` | alive LED, sinks through 1 k from 3V3 | GPIO output, about 1.3 mA | Table 110 (IIO 20 mA per pin) | MATCH |
| 37 | PE7 | TT_ha | `WSEC_A` | voted WiFi changeover, output | GPIO | Table 9 | MATCH |
| 38 | PE8 | TT_ha | `BSEL1` | read-back of voted bank 1, input | GPIO input | Table 9 | MATCH |
| 39 | PE9 | TT_ha | `BSEL2` | read-back, input | GPIO input | Table 9 | MATCH |
| 40 | PE10 | FT_ha | `BSEL3` | read-back, input | GPIO input | Table 9 | MATCH |
| 41 | PE11 | FT_ha | `WIFI_SEC` | read-back of the WiFi changeover, input | GPIO input | Table 9 | MATCH |
| 48, 73 | VCAP | S | `IOCA_VCAP` | LDO output, 2 x 2.2 uF | regulator ON | Table 114 p.211 (CEXT 2.2 uF, ESR under 100 mOhm, two capacitors) | MATCH |
| 51 | PB12 | FT_u | `IOCA_CAN2_RX` | fabric B receive | **FDCAN2_RX, AF9** | Table 10 p.91 (Table 11 p.90) | MATCH; FT_u is supplied by VDD when not in USB use (Table 9 note 7) |
| 52 | PB13 | FT_u | `IOCA_CAN2_TX` | fabric B transmit | **FDCAN2_TX, AF9** | Table 10 p.91 (Table 11 p.90) | MATCH |
| 72 | PA13 | FT | `IOCA_SWDIO` | SWD pads | JTMS-SWDIO, AF0, pull-up after reset | Table 10 p.90 (Table 10 p.89); RM0433 p.533 | MATCH |
| 76 | PA14 | FT | `IOCA_SWCLK` | SWD pads | JTCK-SWCLK, AF0, pull-down after reset | as PA13 | MATCH |
| 81 | PD0 | FT_h | `IOCA_CAN1_RX` | fabric A receive | **FDCAN1_RX, AF9** | Table 10 p.92 (Table 13 p.92) | MATCH |
| 82 | PD1 | FT_h | `IOCA_CAN1_TX` | fabric A transmit | **FDCAN1_TX, AF9** | Table 10 p.92 (Table 13 p.92) | MATCH |
| 92 | PB6 | FT_f | `SCL` | kit bus clock, target | **I2C1_SCL, AF4**, Fm+ capable | Table 10 p.90 (Table 11 p.89) | MATCH |
| 93 | PB7 | FT_fa | `SDA` | kit bus data, target | **I2C1_SDA, AF4** | Table 10 p.90 (Table 11 p.89) | MATCH |
| 94 | BOOT0 | B | `IOCA_BOOT0` | 10 k to GND | boot from BOOT_ADD0, factory 0x0800 0000 (user flash) | RM0433 Table 9 p.138, section 4.4.7 p.181; BOOT0 absolute 9.0 V (Table 109) | MATCH |
| 6 | VBAT | S | `+3V3_IOCA` | tied to the rail | no battery; AN4938: "it is mandatory to connect this pin to an external power supply" | AN4938 Rev 7 section 2.2 p.12 | MATCH |
| 20, 21 | VREF+, VDDA | S | `+3V3_IOCA` | tied to the rail | VDDA 0 to 3.6 V when ADC, DAC, OPAMP, COMP and VREFBUF are unused (Table 112) | Table 112 p.209 | MATCH; AN4938's 100 nF + 1 uF on VDDA is W6-F7, fixed in the r8b candidate (G7) |
| 11, 27, 50, 75, 100 | VDD | S | `+3V3_IOCA` | 3.3 V from a private AP2112K | 1.71 to 3.6 V on LQFP100 (no PDR_ON pin; Table 2 note 5) | Table 112; Table 2 p.22 | MATCH |

## 4. Electrical features the design relies on

| Feature | What the design relies on | H743 (DS12110 Rev 11, revision V section) | Same in Rev 10 and in the revision Y section | H753 (DS12117 Rev 9) | Verdict |
|---|---|---|---|---|---|
| Inputs from rails other than the controller's own (HB1..3 pulled to `+3V3_DEV`, voter read-backs on `+3V3_DEV`, `EMCON_HW` from board C's buffer) | VIN within the operating limit while powered | TT_xx: -0.3 to VDD + 0.3 V; others: up to Min(VDD, VDDA, VDD33USB) + 3.6 V (Table 112 p.209). `+3V3_DEV` (AP63203) and the private rail (AP2112K-3.3) are both nominal 3.3 V; the worst difference of the two regulators' stated tolerances has to stay inside 0.3 V | yes (Table 24 / Table 122) | same | MATCH; the regulator tolerance comparison belongs to the power review (R-PWR) and is not re-derived here |
| A dark controller (LDO held off by `J_IOCOFF_x`, IOHA A4 and A6) with its TT inputs at 3.3 V | no damage and no back-feed | "Input voltage on TT_xx pins" absolute maximum 4.0 V, not VDD-relative (Table 109 p.207); note 3 of Table 110: "Positive injection is not possible on these I/Os and does not occur for input voltages lower than the specified maximum value" | yes: Rev 10 Tables 21, 22 (rev Y) and 119, 120 (rev V) | same | MATCH, and silicon revision V or X avoids erratum 2.2.14 (F1) [revision V only is fitted: SESSION L9T5-D11, record l9t5] |
| FT pins on the kit bus while a controller is dark | the bus is not loaded by a dark controller | FT_xxx absolute maximum Min(Min(VDD..) + 4.0, 6 V), so 4.0 V at VDD = 0, and no positive injection (Tables 109, 110) | yes | same | MATCH |
| Pull-down strength on the 21 controller outputs (100 k today, 10 k owed by FAB-04) | a dark or resetting controller presents high impedance | "During and just after reset, the alternate functions are not active and most of the I/O ports are configured in analog mode" (RM0433 Rev 8 p.533); TT_xx and FT_xx leakage +-250 nA, FT_u +-350 nA (Table 147 p.241) | yes (Table 60 / Table 157) | same | MATCH; the value is FAB-04's, not this page's |
| Supply range and brownout | runs from a 3.3 V LDO; resets cleanly as it falls | 1.71 to 3.6 V on LQFP100; BOR thresholds: VBOR0 1.58 to 1.68 V falling, VBOR3 2.54 to 2.68 V falling, PVD levels to 2.94 V (Table 116 p.212) | yes | same | MATCH; BOR level is a provisioning choice (HC6-SC-5) |
| Output drive | LED at about 1.3 mA; voter inputs (CMOS) | 20 mA per pin, 140 mA total (Table 110) | yes | same | MATCH |
| Thermal grade | inside air 51 C worst | TA to +85 C (suffix 6), TJ to +125 C | yes | same | INSIDE |
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

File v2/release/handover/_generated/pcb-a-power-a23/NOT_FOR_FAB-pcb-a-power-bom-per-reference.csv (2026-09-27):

Reference | Value | Footprint | LCSC | Description | Datasheet | DNP
C1 | 47u 25V | Capacitor_SMD:C_1206_3216Metric
C2 | 47u 25V | Capacitor_SMD:C_1206_3216Metric
C3 | 10u 25V 1210 | Capacitor_SMD:C_1210_3225Metric
C4 | 1u | Capacitor_SMD:C_0603_1608Metric
C5 | 220n | Capacitor_SMD:C_0603_1608Metric | C160828
C6 | 680p | Capacitor_SMD:C_0603_1608Metric | C30816
C7 | 4.7u | Capacitor_SMD:C_0805_2012Metric | C354262
C8 | 4.7u | Capacitor_SMD:C_0805_2012Metric
C9 | 100n 25V | Capacitor_SMD:C_0603_1608Metric
C10 | 100n 25V | Capacitor_SMD:C_0603_1608Metric
C11 | 10u 100V X7R 1210 | Capacitor_SMD:C_1210_3225Metric
C12 | 10u 100V X7R 1210 | Capacitor_SMD:C_1210_3225Metric
C13 | 10u 50V X7R 1210 | Capacitor_SMD:C_1210_3225Metric
C14 | 10u 50V X7R 1210 | Capacitor_SMD:C_1210_3225Metric
C15 | 10u 50V X7R 1210 | Capacitor_SMD:C_1210_3225Metric
C16 | 100n 25V | Capacitor_SMD:C_0603_1608Metric
C17 | 100n 25V | Capacitor_SMD:C_0603_1608Metric
C18 | 3.3u | Capacitor_SMD:C_0805_2012Metric
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

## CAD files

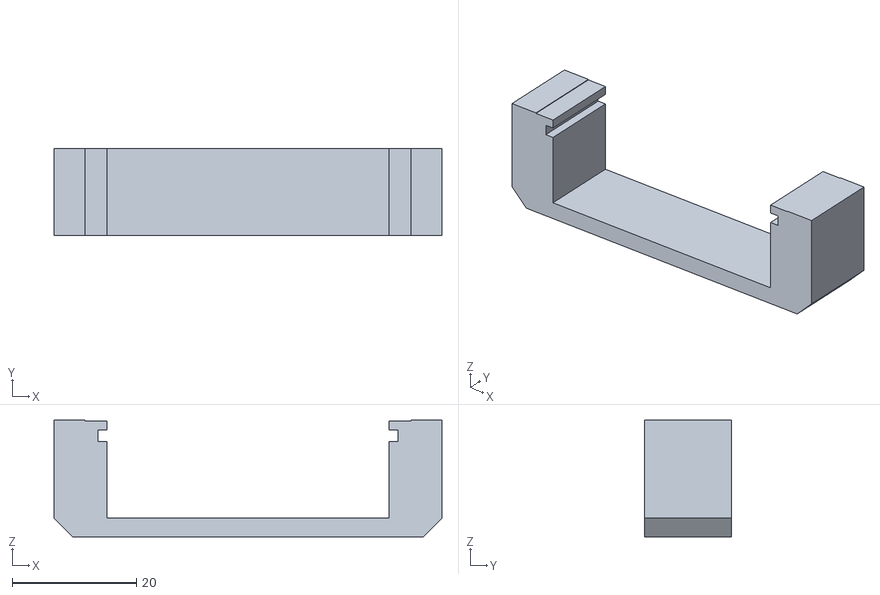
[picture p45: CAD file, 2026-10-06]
compact/v2/coupons/meshsat-coupon_rails.stl
62.5 x 14.0 x 18.8

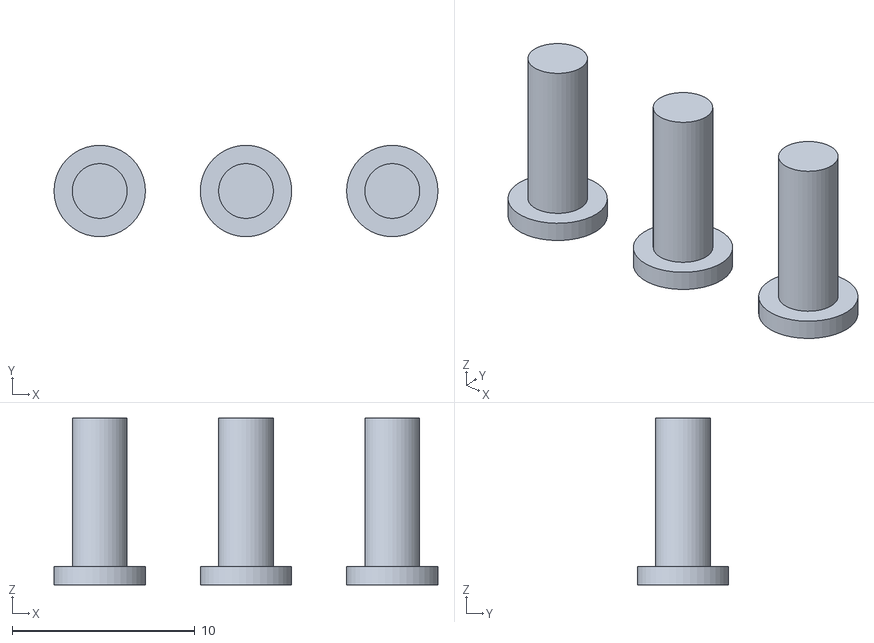
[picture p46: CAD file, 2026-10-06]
compact/v2/print-stl/meshsat-plungers.stl
21.0 x 5.00 x 9.13

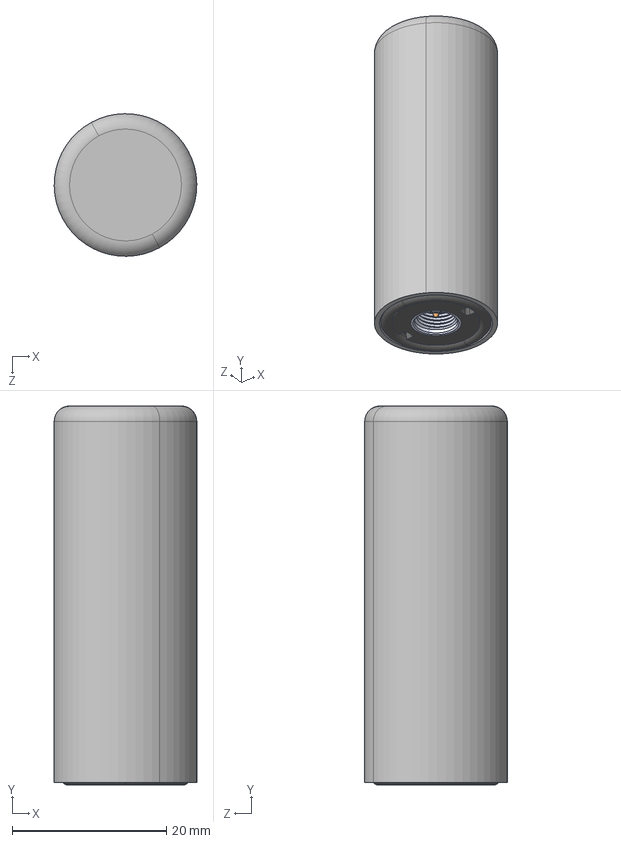
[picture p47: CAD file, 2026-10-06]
compact/v2/reference-cad/groundcontrol-rockblock-9704/Maxtena-helical-antenna-100-00003-02_RevB.STEP
18.5 x 49.2 x 18.5 mm
241-00003-05_View 1
178-00001-01_4.90mm LG x 4

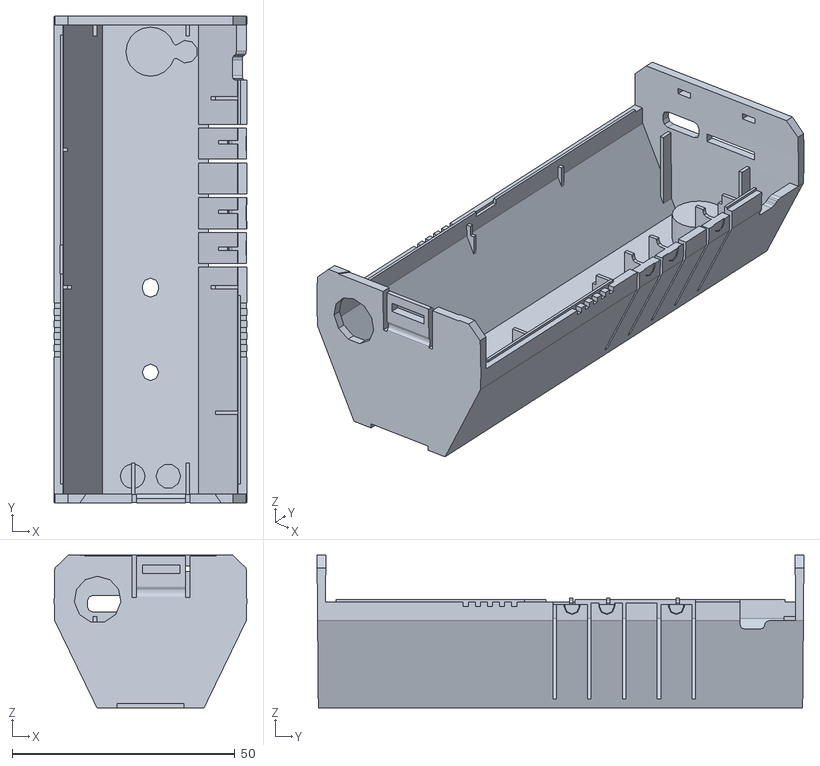
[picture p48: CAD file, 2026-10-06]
compact/v2/reference-cad/lilygo-t-beam-supreme/lilygo-shell/backshell.stl
43.2 x 109.2 x 34.3

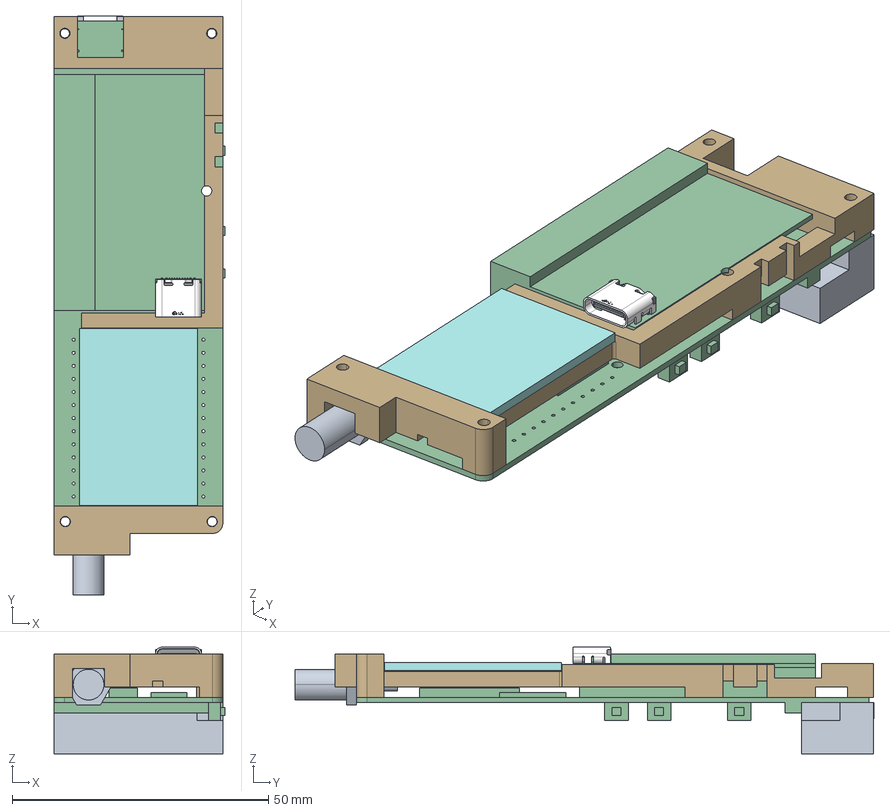
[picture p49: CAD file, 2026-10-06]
compact/v2/reference-cad/lilygo-t-beam-supreme/T-Beam-Supreme-board.stp
33.3 x 112.9 x 20.8 mm
0-PCB_16_1
0-PMMA_59_1
0-TP_7_1
0-TX_4_1
PRT0001_5_1
PRT0001

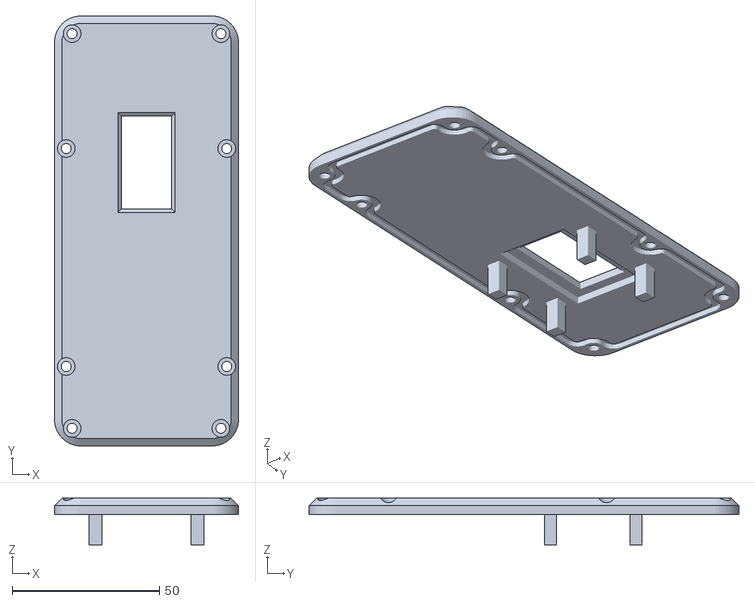
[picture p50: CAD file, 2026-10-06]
compact/v2/validation/build/a_lid.stl
62.5 x 146.0 x 15.8

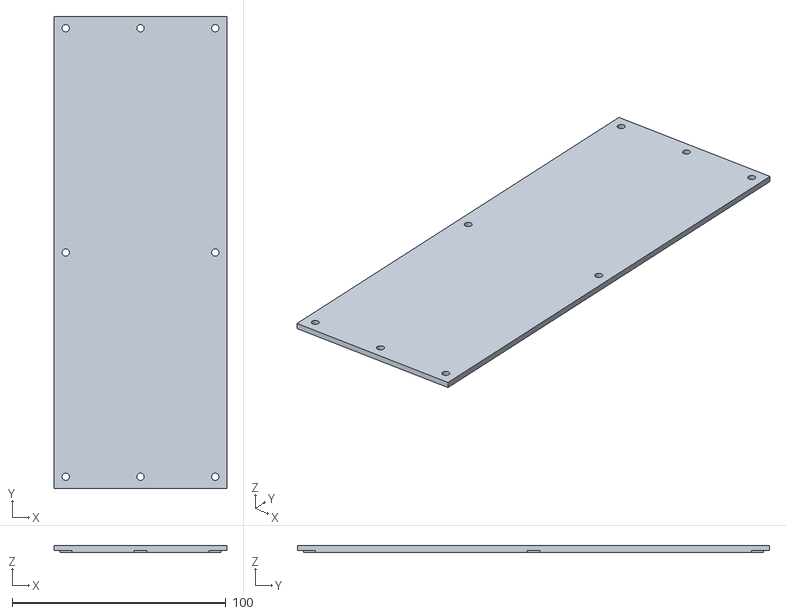
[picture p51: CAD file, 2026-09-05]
v2/cad/render/stl/module_lid.stl
81.0 x 221.0 x 3.50

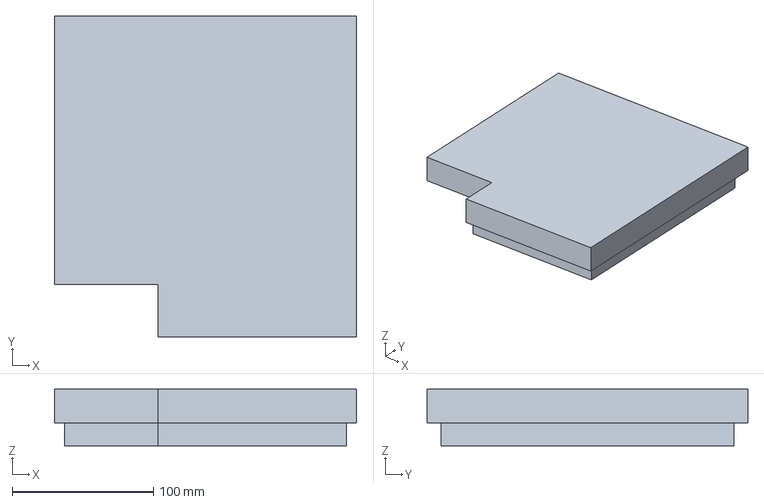
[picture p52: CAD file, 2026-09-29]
v2/docs/records/a1mech/cad/lid-pack-a1-B-envelope.step
213.8 x 227.1 x 40.1 mm

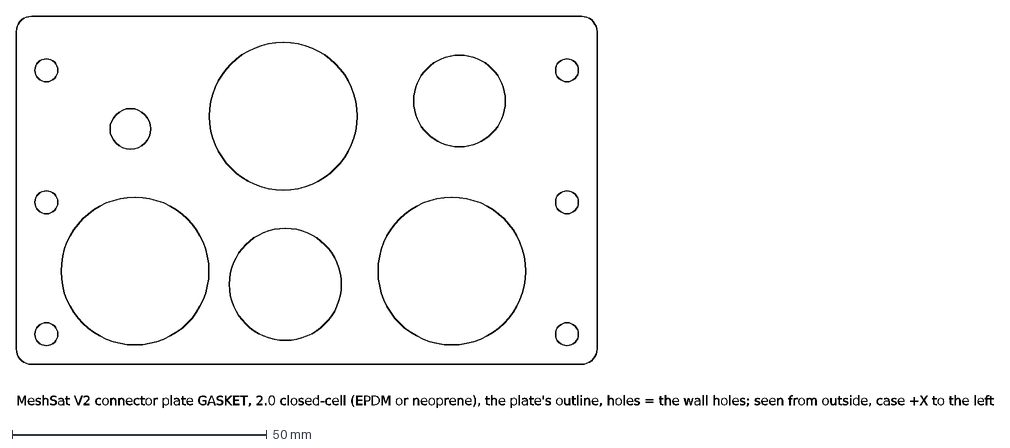
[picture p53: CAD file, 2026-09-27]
v2/release/case-2026-09-27/connector-plate/connector-plate-gasket.dxf
MeshSat V2 connector plate GASKET, 2.0 closed-cell (EPDM or neoprene), the plate's outline, holes = the wall holes; seen from outside, case +X to the left

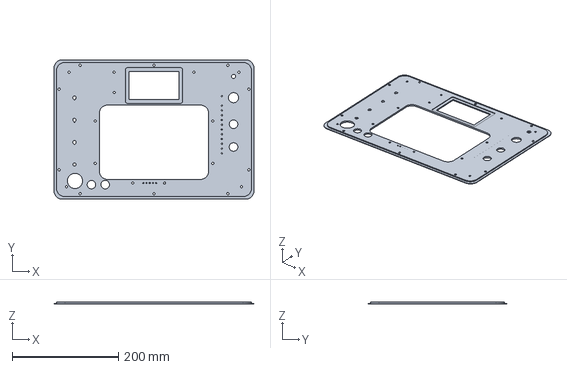
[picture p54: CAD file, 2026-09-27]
v2/release/case-2026-09-27/face-plate/face-plate.step
377.2 x 263.0 x 3.00 mm

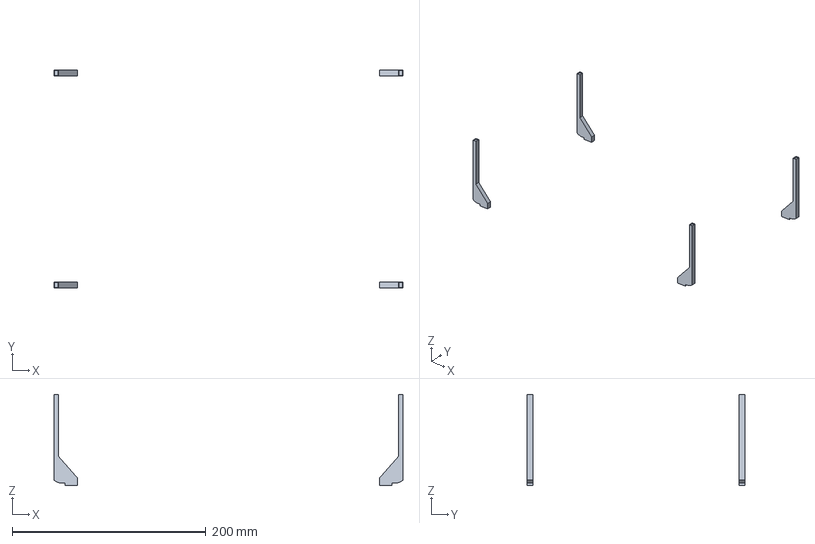
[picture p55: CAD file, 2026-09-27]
v2/release/case-2026-09-27/frame-legs/frame-legs-4.step
360.3 x 224.8 x 94.1 mm

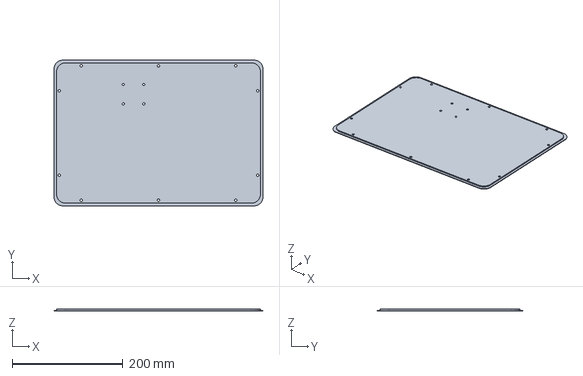
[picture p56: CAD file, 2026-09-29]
v2/release/case-2026-09-27/h1-heat-test-plate/h1-heat-test-plate.step
377.2 x 263.0 x 3.00 mm

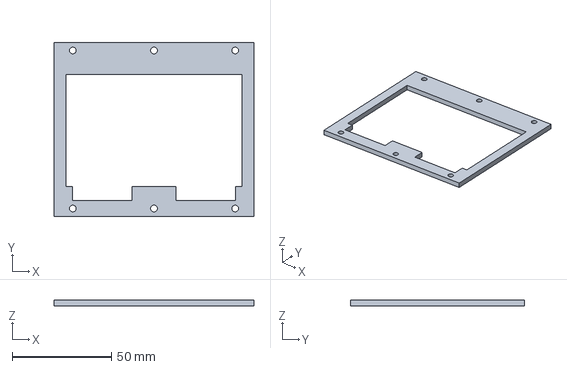
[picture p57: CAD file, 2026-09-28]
v2/release/case-2026-09-27/lid-tray-qmx-r2/lid-tray-qmx-r2-frame.step
101.0 x 87.8 x 3.00 mm

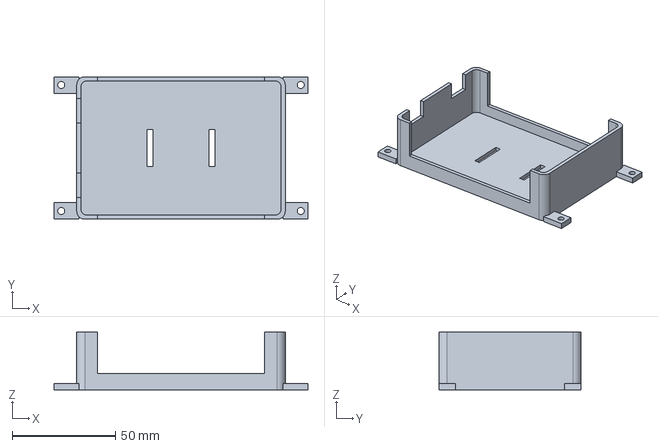
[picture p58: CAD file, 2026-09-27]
v2/release/case-2026-09-27/lid-tray-qmx/lid-bracket-qmx.step
123.0 x 69.0 x 28.0 mm

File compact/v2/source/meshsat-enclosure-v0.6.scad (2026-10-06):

// =====================================================================
// MeshSat stacked enclosure v0.6 - LilyGO T-Beam Supreme over RockBLOCK 9704-SMA
// Units: mm.  Generator: OpenSCAD 2021.01.
//
// v0.6 = response to the 5 Oct 2026 engineering audit of v0.5 (F01-F15).
// Board geometry is registered to the manufacturers' STEP files
// (reference-cad/meshes/*.stl are tessellations of those STEPs) and every
// printed part is clash-checked against them by validation/clash_check.py.
//
// Layout: 9704 (component side down) on edge rails in the lower bay, printed
// separator, Supreme + 18650 in the upper bay, OLED window in the lid.
//
// PART = "assembly"      : printed parts + real board meshes (preview only)
//        "exploded"      : exploded view with ruler + 2 EUR coin
//        "body" "lid" "separator" "membrane" "plungers" "retainer"
//        "molle" "belt"  : printable parts, exported in PRINT orientation
//        "coupon_rimlid" : body top band (grounded) + full lid: gasket/insert/screw coupon
//        "coupon_board"  : upper-bay band with ledges/buttons/window datum (grounded):
//                          drop the separator + real Supreme in, close with the lid
//        "coupon_rails"  : 9704 rail pair + floor strip: real-PCB slot fit coupon
//        "a_*"           : same parts in ASSEMBLED position (for clash checks)
// =====================================================================

PART = "assembly";
$fn = 40;
REF = "../reference-cad/meshes/";       // STEP tessellations (assembly / exploded views)

// ---------------- shell ----------------
wall    = 5.0;
floor_t = 3.0;
lid_t   = 5.5;
cr_out  = 9.0;      // vertical-edge radius
r_bot   = 3.0;      // bottom-edge 45 deg chamfer (bed-facing: chamfer, not fillet - F09)
r_top   = 2.5;      // lid top-edge 45 deg chamfer (lid prints face down; F01: <= lid_t/2)
case_rgb = "#FF6A13";

// ---------------- T-Beam Supreme (LilyGO 3d_file-1105.stp) ----------------
// STEP frame: PCB underside z=0, PCB 1.0 thick, footprint x +/-16.44, y -50..50,
// SMA end at y=-50. Placed rotated 180 deg about Z (SMA end toward the antenna wall).
sup_w   = 32.88;    sup_l = 100.0;    pcb_t = 1.0;
top_max = 10.81;    // tallest top-side part above PCB underside (STEP)
usb_out = 0.95;     // USB-end protrusion beyond PCB edge (STEP: USB-C to y=50.95)
// Battery: holder is not in the STEP. LilyGO's own Supreme shell (same frame) puts the
// holder bottom 18.7 below the PCB underside and its inner roof 0.9 above top_max.
hold_drop = 18.7;   // PCB underside -> holder bottom (LilyGO shell)          [VERIFY]
hold_r    = 10.7;   // holder radius: loose saddles (+2.5 clearance), not a datum [VERIFY]
foam_c    = 1.0;    // compressed thickness of 1.5 mm closed-cell foam under the holder
pad_c     = 1.0;    // compressed thickness of 1.5 mm foam/TPU pads on lid bosses
// PCB retention only where BOTH faces are bare in the STEP: 1.3 mm edge strip,
// board-y 5.7..39.7 from the SMA end, both long edges (validation/heightmap).
edge_strip = 1.3;
seat_by    = [8, 24, 37];      // lower seats (board-y from SMA end)
boss_by    = [8, 37];          // lid hold-downs, directly over seats
sma_clear  = 22.0;  usb_clear = 14.0;
// OLED window: centre matches LilyGO's own shell window within 0.2 mm
oled_cy = 22.75;  win_x = 17.0;  win_y = 31.5;
pane_x = 24.0; pane_y = 38.0; pane_t = 2.0;   // 2.0 mm polycarbonate, exact
pane_clr = 0.3;     // XY clearance per side
bond_t   = 0.2;     // adhesive bond line under the pane
// Side buttons (STEP actuator faces): board-y, depth below PCB underside, protrusion
btn_by    = [50.72, 59.02, 74.65];   // RST, POWER, BOOT
btn_drop  = 1.75;
btn_prot  = 0.38;   // actuator face beyond PCB edge
sup_sma_dx = 9.75;  sup_usb_dx = 7.45;   // offsets from board centreline (case frame)

// ---------------- RockBLOCK 9704-SMA (Ground Control STEP 2A) ----------------
// PCB 47.8 x 52.0 x 1.5, component side DOWN: module +5.9 on top; supercaps,
// SMA, header pins, USB-C below (to -10.3 / SMA -11.1). Edges bare within 1.45 mm.
rb_w = 47.8;  rb_l = 52.0;  rb_pcb = 1.5;  rb_h = 5.9;
rb_lift   = 12.5;   // PCB underside above floor (lowest part 1.4 mm off floor)
rb_slot   = 1.80;   // FDM slot height (GC moulded mount: 1.70 +/-0.05). Tune with coupon_rails.
rb_engage = 1.2;    // lip engagement on each PCB edge
rb_sidec  = 0.3;    // side clearance
rb_sma_dx = 8.45;  rb_sma_z = -6.35;  rb_sma_out = 7.2;

// ---------------- derived cavity ----------------
in_w   = 52.5;
in_l   = sma_clear + sup_l + usb_clear;            // 136.0
ledge_z = rb_lift + rb_h + 0.8;                    // separator underside
sep_t  = 3.0;
sup_z0 = ledge_z + sep_t;                          // separator top
pcb_z  = sup_z0 + foam_c + hold_drop;              // Supreme PCB underside
in_h   = pcb_z + top_max + 1.5;                    // 1.5 mm over the tallest part
body_h = floor_t + in_h;
out_w = in_w + 2*wall;  out_l = in_l + 2*wall;
cx     = in_w/2;                                   // board centreline (both boards)
sup_x0 = cx - sup_w/2;
sup_ytop = in_l - sma_clear;                       // Supreme PCB SMA-end edge
function by(b) = sup_ytop - b;                     // board-y -> cavity y
rb_x0 = cx - rb_w/2;
rb_y1 = in_l - sma_clear;   rb_y0 = rb_y1 - rb_l;

// ---------------- screws / seal ----------------
pil_r = 7.0;  insert_d = 4.0;  insert_h = 7.0;     // M3 heat-set, <=5.7 long: pocket 7.0
screw_d = 3.4; head_d = 6.0; head_h = 3.2;        // lid: M3x8 -> 5.7 below mating face
cord_d  = 2.0;                                     // F07: 2.0 mm silicone cord
g_in = 1.15; g_out = 3.85; groove_d = 1.5;         // 2.7 x 1.5 -> 77.6 % fill, 25 % squeeze
mid_ys  = [22, in_l - 40];
pillars = concat([[1,1],[in_w-1,1],[1,in_l-1],[in_w-1,in_l-1]],
                 [for(y=mid_ys) [-1,y]], [for(y=mid_ys) [in_w+1,y]]);
function is_corner(p) = (p[1] < 5 || p[1] > in_l-5);

// ---------------- ports ----------------
sma_hole = 6.6;
lora_bh  = [39, pcb_z + 3.5];          // x,z on the top wall
iri_bh   = [14, 9];
usbc_hole = 16.2;   usb_bh = [18, 10.5];  // [VERIFY] against the chosen panel USB-C (nut up to 20 mm OD)
vent_d    = 12.3;   vent_by = 35;  vent_z = 9;   // vent on the RIGHT side wall, lower bay
// SOS (12 mm IP67 momentary), guarded; switch body must stay below the Supreme
// SMA-end overhang (STEP: z >= PCB underside + 1 out to board-y -4.2)
sos_hole = 12.2;  sos_depth = 20;  sos_x = 17;  sos_z = pcb_z - 6.5;
shroud_id = 21;  shroud_od = 27;  shroud_h = 8;  drain_w = 3;  drain_h = 1.5;

// ---------------- carry plates ----------------
rear_ins_h = 7.0;
plate_t = 3.0;
strap_w = 26.5;  strap_gap = 3.6;  molle_pitch = 38.1;  skin_t = 2.4;  rail_t = 2.5;
belt_w = 40;  belt_gap = 5.6;
tab_l = 14;  lanyard_slot = [16,6];
rear_pts = [[wall+1,wall+1],[out_w-wall-1,wall+1],[wall+1,out_l-wall-1],[out_w-wall-1,out_l-wall-1]];

// ---------------- side buttons: membrane + guided plungers ----------------
btn_y     = [for(b=btn_by) by(b)];          // cavity y
btn_z     = pcb_z - btn_drop;               // cavity z
btn_face  = sup_x0 - btn_prot;              // actuator face, cavity x
pl_gap    = 0.3;                            // plunger-to-actuator gap at rest (no preload)
pl_travel = 0.65;                           // hard stop: max plunger travel
strip_y0  = min(btn_y) - 8;  strip_len = max(btn_y) - min(btn_y) + 16;
flange_t = 1.5;  pocket_d = 1.2;            // 0.3 mm (20 %) flange compression, wall is the stop
fl_h  = 14;      ret_t = 3.0;  ret_h = 24;  // retainer covers flange + screw rows
cap_d = 5.4;     cap_out = 0.8;             // cap protrudes 0.8 mm
pl_head_d = 5.0; pl_head_t = 1.0; pl_d = 3.0;
ret_screw_dy = [3, strip_len/2, strip_len-3];   // 6x M2x6: rows at +/-9.5 mm

assert(r_top <= lid_t/2, "lid round-over would breach the mating plane");
assert(groove_d < lid_t - r_top, "groove too deep for lid");
assert(sos_z + sos_hole/2 + 0.3 < pcb_z + 1, "SOS switch would hit the Supreme SMA-end overhang");

// =====================================================================
module rbox(w,l,h,r){ linear_extrude(h) offset(r) offset(delta=-r) square([w,l]); }
// slab with rounded vertical edges (rv) and 45 deg chamfers on the bottom (rb) / top (rt)
// edges; clipped to 0..h so no edge treatment can cross a mating plane (F01)
module rshell(w,l,h,rv,rb,rt){
  intersection(){
    hull() for(x=[rv,w-rv], y=[rv,l-rv]) translate([x,y,0]) rotate_extrude($fn=56)
      polygon([[0,0],[rv-rb,0],[rv,rb],[rv,h-rt],[rv-rt,h],[0,h]]);
    translate([-1,-1,0]) cube([w+2,l+2,h]);
  }
}
module at_in(){ translate([wall,wall,floor_t]) children(); }
module cavity2d(){
  difference(){ offset(r=1.5) offset(delta=-1.5) square([in_w,in_l]);
                for(p=pillars) translate(p) circle(pil_r); }
}
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

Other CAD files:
compact/v2/reference-cad/meshes/supreme_step.stl
v2/release/case-2026-09-27/rf-entry-plates/rf-entry-gasket-west.dxf
v2/release/handover/H1/v2/release/revA/case/lid-bracket-qmx/lid-bracket-qmx.step
v2/release/handover/H1/v2/release/revA/case/pack-4s/pack-4s-lid.step
compact/v2/coupons/meshsat-coupon_board.stl
compact/v2/coupons/meshsat-coupon_rimlid.stl
compact/v2/print-stl/meshsat-belt.stl
compact/v2/print-stl/meshsat-body.stl
compact/v2/print-stl/meshsat-lid.stl
compact/v2/print-stl/meshsat-membrane.stl
compact/v2/print-stl/meshsat-molle.stl
compact/v2/print-stl/meshsat-retainer.stl
compact/v2/print-stl/meshsat-separator.stl
compact/v2/reference-cad/groundcontrol-rockblock-9704/Mount_for_RockBLOCK_9704-SMA_RevA.STEP
compact/v2/reference-cad/lilygo-t-beam-supreme/T-BEAM-SUPREME-V3.0.DXF
compact/v2/reference-cad/lilygo-t-beam-supreme/lilygo-shell/brackets.stl
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

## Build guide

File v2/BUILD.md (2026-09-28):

# Building a V2 kit from this repository

**Status (27 September 2026): the build guide of the 7 September generation, kept as history and as the one end-to-end
account of how a kit goes together. Do not order boards from it.** No board of the set is ready for layout
(`docs/CURRENT-EVIDENCE.md`: "Foundations incomplete; 0 boards ready for layout; 0 physically verified"); every
deliverable folder predates the circuit corrections of 26 September 2026 (`faf8c981`, `458b2873`, `d90f30e4`) and
every later one, which are in the schematics only; and the order folder `release/revA/order/` is rebuilt and quarantined, with nothing
ordered from it (owner decision 41 of 25 September 2026). The lines of this page that contradicted the current
baseline are corrected in place and marked "(corrected 27 September 2026)". Where this page and `docs/CASE-MARGINS.md`
section 4, `docs/PANEL.md`, `docs/CONOPS.md` or `docs/V2-SPEC.md` still differ, those documents govern. Keeping the
page as history with its stale lines corrected, rather than withdrawing it, is the session's choice SC-15 under the
owner's standing rule of 26 September 2026: it is the only assembly narrative in the tree, and the head above keeps a
reader from ordering from it. Reverse by withdrawing the page or its section 1.

The MESHSAT-830 generation of the carrier set (7 Sep 2026) has been designed and generated; no board of it has been fabricated and no kit has been built. This page was written as the path from an empty JLCPCB cart to an assembled kit, in order, pointing at the documents that carry the detail. Read it together with `docs/ASSEMBLY.md` (fasteners, build order, the pack, leads, coating, labels, removal, bench checks, bench-fit lists), `docs/PANEL.md` (the panel controller contract), `docs/V2-SPEC.md` (the device set and the budgets) and `docs/TEST-PLAN.md` (the qualification plan). The design record with every number and every ruling is `docs/MESHSAT-709-geometry-appendix.md`; sections 32.49 to 32.61 are this generation.

MeshSat is a prototype. Expect changes after the first build.

## 0. Before you start

- The rulings that are not open for redesign (appendix 32.49 to 32.53): three identical Compute Module 5 slots on one carrier, most radios and the sensor and panel controllers USB devices shared by the HAL, k3s across the three modules (corrected 27 September 2026: not every device is a USB device; the LoRa module is on slot 3's SPI, the 5G module's data on slot 2's PCIe lane, the two WiFi link cards on the PCIe switches of slots 1 and 3, and the compute modules' own radios on the modules, `docs/V2-SPEC.md` correction 6; the LoRa module and cellular data are the named exceptions to the failover requirement for prototype 1, session choice SC-02); a built 4S smart pack in the east pocket (appendix 32.62; the BB-2590/U of 32.49 did not fit the case) with the charger, gauge reading and power control on PCB-A; no vent opening anywhere in the case, the plate or the connector plate (internal IP68-rated fans carry the heat to the skin); EMCON is a hardware line from the panel toggle, plus a software hold, meant to silence every transmitter (corrected 27 September 2026: as generated the line is drawn to every transmitter, but none is yet dark end to end; the radio's own chain closes at desk for 15 of the 17 and is open for the SA868, whose PTT threshold is unpublished, and the RockBLOCK 9704, which runs on its own supercapacitors with its ENABLE held by firmware once its supply is cut, the 5G module's supply being removed by hardware at once since board B's round 8 (SD-EMC-1r8); every row also waits on the shared items and the session's latency limit, and none has been shown on a bench, `docs/feasibility/EMCON.md` section 0a, feasibility blocker FEA-002); the panel is a USB device driven per `docs/PANEL.md`.
- Nothing is to be ordered from this page (corrected 27 September 2026). The document check of every COTS site against the manufacturer's own drawing (appendix 32.1; the documents are in `vendor/`, rows marked "previous generation" belong to the released set of 5 and 6 September) was the gate of 7 September. What gates a board today is its layout entry and then its fabrication release (`docs/EXECUTION-PLAN.md`, stage gates; the blockers per board in `docs/CURRENT-EVIDENCE.md`), and the order folder is quarantined (decision 41).
- The software of this generation is specified but not written: the panel controller firmware (MESHSAT-837), the sensor controller (838), the HAL device sharing and the per-device services (835 to 848). Corrected 27 September 2026: until the panel controller's firmware drives them, board A's slot enables stay low and no compute module runs (`docs/PANEL.md` section 7; adjudication A01, `docs/records/adj/`); the panel, the radios and the sensors come alive with that software.

## 1. The boards (not for ordering)

Corrected 27 September 2026: this section was "Order the boards". The order folder `release/revA/order/` was rebuilt from the deliverable folders and quarantined on 25 September 2026 (owner decision 41, appendix 32.365); each `ORDER-NOTES.txt` opens with its board's readiness, and every board reads NOT_READY (`release/revA/order/README.md`). No cart line is touched and nothing is ordered. The folders, with the phase each holds against the phase its board declares:

| Board | Folder in `release/revA/order/` | Folder phase | Declared phase | Size (mm) | Layers as generated |
|---|---|---|---|---|---|
| PCB-A POWER + I/O | `PCB-A-POWER-A22/` | A22 | A32 | 240 x 160 | 6, JLC06161H-3313 (In1 and In4 solid ground) |
| PCB-B COMPUTE | `PCB-B-COMPUTE-B16/` | B16 | B21 | 330 x 200 | 6, JLC06161H-3313 (In1 solid ground, In4 the 5 V planes); an eight-layer measurement ruled first (decision 43) |
| PCB-C PANEL BACKER | `PCB-C-DISPLAY-C24/` | C24 | C24 | 344 x 228 ring, 240 x 176 void | 4, JLC04161H-7628; six layers ruled (decision 27), not yet regenerated; the face itself is the aluminium plate of `release/case-2026-09-27/face-plate/` (case choice C1) |
| PCB-D VHF APRS | `PCB-D-APRS-D8/` | D8 | D12 | 100 x 80 | 4, JLC04161H-7628 |
| PCB-E1 DOCK STRIP | `PCB-E1-DOCK-E6/` | E6 | E17 | 267 x 68 | 4, JLC04161H-7628 |
| PCB-E5 DOCK BLOCK | `PCB-E5-BLOCK-E5/` | E5 | E5 | 43 x 26 | 2, standard, 2 oz outer copper |
| PCB-P PACK BMS | `PCB-P-PACK-P4/` | P4 | P4 | 70 x 44 | 2, standard, 2 oz outer copper; four layers at 2 oz ruled (decision 28), not yet regenerated |

No layout of boards A, B, C, D, E or P carries its board's corrected schematic, including C and P, whose folder phase equals the declared phase: SCH-002 reads FAIL on A and B and INCONCLUSIVE on C, D, E and P (`docs/CURRENT-EVIDENCE.md`). E5 has no schematic; its board file is its design.

The settings the 7 September order notes gave, kept for the record: 1.6 mm FR-4, 1 oz outer copper (0.5 oz inner), ENIG, matte black solder mask, white silkscreen, no castellations, order number removed, quantity 5 (the JLCPCB minimum), 90 ohm differential tuning on the USB 2.0 pairs (0.2 mm track, 0.15 mm gap on the outer layers) and, on B, 100 ohm on the PCIe, USB 3 and HDMI pairs (0.127 mm track and gap on the six-layer stack). The fine-pitch parts (the six Compute Module receptacles, the PCIe switches, the USB 3 hubs, the RP2040 on C) took 0.40/0.20 mm vias, 0.127 mm tracks and clearance and a 0.19 mm hole-to-copper clearance, the rules of Raspberry Pi's own CM5 IO board. Both free confirmation options (production file review and the BOM/CPL confirmation) were to be on, and the rotation of every polarised part checked against `release/revA/review/<board>/*-assembly-top.pdf`.

Parts JLCPCB does not fit are listed per board in the ORDER-NOTES ("fitted at the bench") and in `docs/ASSEMBLY.md` section 9: the Compute Modules and their receptacle-mounted cards, the bought modules (RockBLOCK, LimeSDR, the QMX unit, the sensor modules), the PA module, the connectors on flying leads and the switches.

A board is regenerated by its generators (`README.md`, "Regenerating a board"); `make_handoff.py` then rewrites `order/` and `review/`.

## 2. Everything else to buy

Case and face: Peli 1450 without foam and the 1450PF panel frame. Corrected 27 September 2026 (the session's case choices C1 and C6, `docs/CASE-MARGINS.md` section 4): the face plate lies on top of the frame over Peli's o-ring and is screwed from above into Peli's brass inserts with ten 6-32 UNC x 1/2 in A2 pan-head screws, and the frame stands on four setting legs cut from 6.0 mm 6061-T6 plate, bonded under its ring; the plate is 377.2 x 263.0 x 3.0 mm with a rebated band, which the plate generator carries since `c351115d`. The face plate is a CNC part from the DXF and STEP in `release/case-2026-09-27/face-plate/` (5754 or 6061, 3 mm, black anodised, laser-marked from the SVG); the sixteen LEDs need sixteen Mentor 1282.5004 light guides (and the hardware EMCON lamp of board C's round 8 a seventeenth once its hole is in the plate, open item S-44), the backer eight PEM SO-M3-10 standoffs, the PA module two PEM S-M3 nuts pressed into the plate's underside. The QMX lid tray is the r2 set `release/case-2026-09-27/lid-tray-qmx-r2/` (sheets 14r2-1 to 14r2-3; the r1 tray and sheet 14 are superseded): the tray (68 g) and its retaining frame (12 g) printed in Prusament PC Blend at 100 percent infill, a 2.0 mm 5052-H32 lid plate cut from its DXF and bonded to the lid with DP8005, ten M3 x 5 countersunk A2, six M3 x 10 button head A2 with six M3 square nuts, and two PORON 4701-30 pads; the harness's crossing of the sealed face is not designed yet (S-95); the tablet bracket for the west third of the lid is still to be drawn (appendix 32.60 item 5).

The monitor: Xenarc 709GNK (IP67, 7 inch, HDMI and USB touch, 12 V) with its cable set; it sits IN the plate with its glass level with the aluminium, held by a rear frame on four M4 with its connector block through the plate cutout, so the HDMI, USB and 12 V leads run below the plate to B and A.

Modules that mount on the boards (one kit, appendix 32.49): three Raspberry Pi Compute Module 5 (8 GB, 64 GB eMMC, wireless, CM5108064) with three CM5 Coolers, three M.2 2242 NVMe drives (a -20 C or industrial grade, `docs/feasibility/POWER-THERMAL.md` section 9.4), two AsiaRF AW7915-AED M.2 E-key WiFi link cards with their MHF4 pigtails (slots 1 and 3; not rated to the envelope's -20 C, from 0 C in the maker's 2023 PDF and -10 C on its current page, the same section), a Quectel RM520N-GL 5G module in the M.2 key-B socket with its pigtails on ANT0 and ANT2 (and ANT3 under owner ruling D-07) and two nano-SIMs (slot 2; corrected 27 September 2026: the dual SIM is two nano-SIM holders, with an eSIM-plus-nano-SIM build possible with an eSIM-fitted module variant, `docs/V2-SPEC.md` correction 22), a LimeSDR Mini 2.4 in its USB 3 bay (rated from 0 C), a RockBLOCK 9704 with the Ground Control bracket and the Maxtena helical antenna, a Quectel YEGD006U1A GNSS puck, and the Ebyte E22-900M30S LoRa module, the two Ebyte E72-2G4M20S1E radios (Zigbee coordinator and Thread RCP), the Quectel LG290P and the NiceRF SA868 VHF module (fitted by the assembler where JLCPCB has them, else at the bench). The QMX HF transceiver is bought assembled from QRP Labs and rides in the lid tray with its USB-C lead, 12 V lead and BNC-to-SMA jumper; the wire antenna kit and tuner are the operator's. The Pervasive Displays E2370KS0C1 e-paper goes on the backer's 24-way ZIF. The Mitsubishi RA30H1317M1 amplifier module bolts under the plate. Sensor modules on E's headers: a RadiationD-class Geiger counter board with an SBM-20 tube, a DCF77 receiver module, a CJMCU-3935 lightning sensor board, and the outside pod (BME688 and AS7331 on a small board in a sealed housing on the connector plate, over an M8 sealed receptacle; no CAD model of the pod exists in `v2/cad/` yet). A CR2032 for B's holdover clock. A USB camera module of about 25 x 25 mm for the plate's sealed window (part owed). Five IP68 fans (three on the coolers, two mixers on E, JST-SH leads).

Battery (corrected 27 September 2026, owner ruling D-06 of 26 September 2026): one 4S3P block of twelve Samsung INR18650-35E cells, about 145 Wh, shrink-wrapped with no rigid enclosure, in the east pocket under B's overhang, its fit designed against Peli's own figures (`docs/CASE-MARGINS.md`); the BMS board P (the BQ4050 SMBus gauge with protection and balancing, two high-side N-FETs, the 2 mohm shunt, the 25 A blade, the tap, thermistor and SMBus headers; since `faf8c981` and `d90f30e4` its schematic also carries the second-level protector, the chemical fuse and the gauge's PTC input of owner ruling D-15, which no board P layout carries yet); the XT60 lead and the SMBus lead to E. The printed enclosure of `v2/cad/pack_4s.py` fits neither pocket and is to be redesigned around the shrink-wrapped block (a session item under D-06). The RS PRO 245-556 heater mat goes under the block on A's `J_HEAT`, fed a regulated 12 V (`docs/V2-SPEC.md` correction 2). No second pack has a location: owner ruling D-01 defers it (`docs/CONOPS.md` section 2a). The pack is not built before the paid battery-and-protection review of owner ruling D-09 (`docs/review-packets/battery/`).

Solar (optional): a bare 12 V class panel of your choice, up to about 100 W, wired to the spare pair of the shore plug; E's tracker regulates it. No panel part is prescribed.

Hardware per `docs/ASSEMBLY.md` section 1: four M3 stainless rods with Nyloc nuts, spacers for the dock gap and for the A to B bay, four M3 x 22.6 standoffs for the D mezzanine on A, twelve M2.5 x 4 standoffs with screws for the three Compute Modules, M2.5 standoffs for the seven M.2 sockets, four M3 x 6 standoffs for the raised dock block, ten 6-32 UNC x 1/2 in pan heads for the plate (corrected 27 September 2026, C1; was ten M3 x 8 with star washers), four M4 x 8 for the Xenarc, two M3 x 8 for the PA flange, two M3 x 6 for each cooler fan.

Consumables: 3M 467MP or 9495LE transfer tape (the e-paper), 3M VHB 5952 pads (dock strip and the setting legs), MG Chemicals 422B acrylic conformal coating, kapton for the masks, IPA, thermal pad 1.0 mm for the PA flange.

Electrical: the Preci-Dip 813-S1-012-10-016101 spring-loaded connector for A's `J_DOCK` (2 x 6 at 2.54 mm, 7.0 mm high, solder tails), nine Mill-Max 0858 class 9 A spring pins for the pack contacts and the pre-charge pin, eleven blind-mate RF receptacles with their right-angle plugs as generated (twelve with D-07's third 5G jack), Keystone 3568 mini blade holders with a 25 A blade on A (`F1`, the pack node) and a 25 A, two 10 A on E (`F3` pack, `F1` vehicle, `F2` solar), JST-VH leads with 16 AWG for the three slot rails, the device rail, the PA rail, the HF rail, the PoE rail, the monitor and the D mezzanine, JST-XH leads for the MAIN and PI buttons and the heater, JST-PH leads for the two headset jacks, the camera, the QMX USB, the PA gate bias and the wall USB pairs, U.FL and SMA pigtails per the table in `docs/ASSEMBLY.md` section 4, twelve hook-up wires and a 12 AWG pair from the dock strip up to the contact block.

Wall parts (corrected 27 September 2026, the session's case choices C2 to C4, `docs/CASE-MARGINS.md` section 4). On the back wall, one 114 x 68.3 x 5 mm aluminium connector plate between the hinge fairings, outside the wall on a 2 mm closed-cell gasket, on six M4 x 25 with bonded sealing washers, carries: a Glenair D38999 receptacle for the vehicle and shore DC pair plus the solar pair with its D38999/26 plug, size 16 contacts and strain relief, 2 m of 4 x 1.0 cable (Lapp OLFLEX ROBUST 210 or Alpha Wire 25064) and a NATO 2-pin vehicle plug on the vehicle lead; the Glenair 233-370 USB receptacle, which carries the wall data path and is the console and key-fill port (owner ruling D-12); a sealed Gigabit RJ45 receptacle (PoE out), to be picked inside a MIL-DTL-38999 shell 15 envelope, with a voltage rating that covers the 54 V PoE feed; a sealed USB-C receptacle, the 45 W outlet, which carries power only (D-12); the M8 receptacle of the sensor pod; a ground stud. In the end walls, twelve PolyPhaser GTH-SFF-AL gas-discharge arrestors are the antenna bulkheads, at Z 59 on one 6.0 mm aluminium RF entry plate per wall on its gasket (eight M4 x 12 A2 button heads on sealing washers per plate): east, south to north, 5G MAIN, 5G DIV, the third 5G jack of D-07, IRIDIUM, LORA; west VHF, HF, WIFI 2.4, GNSS, SDR, WIFI P2P A, WIFI P2P B. The case generators (`tools/panel1450.py`, `tools/case_wall_cutouts.py`) carry this layout since `c351115d`, with its templates in `release/case-2026-09-27/templates/`; `release/revA/case/wall-receptacles-1to1.pdf` is the superseded 7 September layout (eleven Amphenol Connex 132170 couplers in 6.5 mm D-holes at Z 88 and a 54 x 82 plate between the ribs), kept as history.

Panel hardware: SW_MAIN C&K ATP19-SL1-603-B0SA-03G (19 mm, green ring), SW_PI C&K ATP16-SL1-403-M0SA-04G (16 mm, amber), SW_TEST C&K ATP16-SL1-203-M0SA-04G (16 mm, white), the LIGHTING toggle NKK M2044SD3A01 on its D3 splashproof bushing with the AT428H boot, three APEM 5636ADKB-2V locking toggles (SW_SOS, SW_EMCON, SW_ZERO; hinged safety covers on SOS and ZEROIZE, cover part owed), the Floyd Bell MC-09-530-Q IP68 sounder with its 61663 gasket, two U-174/U headset jacks (Amphenol Nexus class, drawing owed), the sixteen 3 mm LEDs of the backer. Panel seals: 1.0 mm Silex GP60 silicone sheet for the bezel washers, a 2.0 mm UV-grade polycarbonate lens over the e-paper window on 3M VHB 5915 with 3M Primer 94, DOWSIL 3145 clear silicone; Peli's own o-ring under the plate (corrected 27 September 2026, C1: the PORON 4701-30 frame gasket ring is dropped); Glenair 930-001 flange gaskets and bonded washers for the connector plate; a 3M 7871EC polyester label for the serial number.

## 3. Prepare the case

1. Corrected 27 September 2026 (C6): bond the four setting legs under the 1450PF frame's ring with the printed corner locators, lower the frame on its legs into the case, centre it, and fix it with Peli's four screws as Peli instructs; Peli's ten inserts are the face plate's screw pattern (`release/case-2026-09-27/drawings/`, sheet 1 the face plate and sheet 2 the frame and legs).
2. End walls (corrected 27 September 2026, C2 and C4): cut the 27 mm holes at Z 59 (five on the east wall, seven on the west) and eight 5.0 mm screw holes per wall; fit the arrestors on each RF entry plate on the bench, then each plate on its gasket from outside with its eight M4 x 12. The east and west wall templates are in `release/case-2026-09-27/templates/case-templates-1to1.pdf`, from `case_wall_cutouts.py`, which carries C2 since `c351115d`; sheets 3 and 4 of `release/revA/case/` show the superseded eleven 6.5 mm D-holes at Z 88.
3. Back wall (corrected 27 September 2026, C3): the connector plate centred at X 0, Z 18.3 to 86.6, outside the wall between the hinge fairings, over three 29 mm, one 22, one 18 and one 8 mm wall holes and six 4.5 mm screw holes; fit the plate with its gasket, the two Glenair receptacles, the RJ45, the USB-C, the M8 pod receptacle and the ground stud; the sensor pod screws onto the plate over the M8. The back-wall template is in the same file; sheet 1 of `release/revA/case/` shows the superseded window between the ribs at X -95 and -18.
4. Dock strip E on the floor along the front wall: degrease with IPA, four VHB pads at the corners, locate it by dropping two rods through its south rod holes before the pads touch.
5. The pack in the east pocket (corrected 27 September 2026, D-06: the block's west face at X 122, centred in Y, `docs/CASE-MARGINS.md` section 4) with the heater mat under it.
6. Bulkhead legend strips beside the arrestor rows (the west and east lists above), the "RF HAZARD DURING TX" label next to the VHF arrestor, the asset label in Peli's recess (`docs/ASSEMBLY.md` section 6).

## 4. The pack

Corrected 27 September 2026: the pack is built for the kit (appendix 32.62) as one 4S3P block of Samsung INR18650-35E cells welded on nickel strip and shrink-wrapped (owner ruling D-06), with the BMS board P and its SMBus gauge, protection and cell thermistors, and it lies in the east pocket. It is not built before the paid battery-and-protection review of D-09. Its XT60 lead plugs into E's `J_BATT` (pin 2, the pad nearer `F3`, is positive) and its SMBus pair into `J_SMB`. A's BQ25731 charger (SMBus 0x6B) charges it from the 9 to 36 V front end; the charger has no conductor to the pack's gauge, which the sensor controller on E reads (corrected 27 September 2026, `docs/PANEL.md`, item 3 of the note at its head; adjudication A07), so the battery bar on the panel is the pack's state of charge as the sensor controller reports it. The pack is fused at 25 A on E (`F3`) and again at A's node (`F1`), and board P's schematic carries the second level of D-15 (not yet laid out). Charge current and the JEITA window are the charger's settings. The pack's own qualification (shock, vibration, temperature) is part of the kit's programme in `docs/TEST-PLAN.md`; the gauge takes its golden image from TI's bqStudio on the bench before the pack is closed.

## 5. Assemble

Follow `docs/ASSEMBLY.md` section 2 step by step; the short form, as of 7 September (board names by letter; the fitted boards are those each folder of section 1 holds):

1. Dock strip E: solder the leads (`J_DCIN`, `J_SOLAR`, `J_BATT`, `J_SMB`, the sensor headers, the two mixer fans), fit the three fuse holders with their blades, and check the front end gives the 20 V bus at the block lands with 9 V and 36 V in. Then fit the raised block E5 on its four 6 mm standoffs, solder the twelve signal wires and the 12 AWG pair from the strip into the block's plated lands from below, and stick the strip down on its VHB pads.
2. Rods through the strip's holes with the spacers that set the dock gap (washer stack under the two north rods so all four sit level).
3. PCB-A: solder the Preci-Dip connector and the nine Mill-Max pins in from the underside (tails on the top face), fit the blind-mate receptacles, the 25 A blade, and lower the board onto the rods so its pins land on the block; check continuity from the block's lands to the board with a meter before the first power-up.
4. PCB-D on A's four 22.6 mm standoffs at the mezzanine site: the 2x8 harness ribbon into `J_MEZZ1`/`J_HARN1`, the 5 V lead into `J_PWR1`, the antenna pigtail from `J_ANT` to A's VHF jack `J_RF1`; the PA drive coax (`J_PAIN`), the PA output coax (`J_PAOUT`), the gate bias lead (`J_VGG`) and A's 13.8 V lead (`J_PA`) are left coiled for the plate.
5. Bay spacers, PCB-B: the three Compute Modules pressed onto their receptacle pairs and screwed to the standoffs, the coolers clipped on with their fan leads in `J_FAN1..3`, the NVMe drives in `J_M2N1..3`, the WiFi link cards in slots 1 and 3 with their pigtails to the WIFI P2P entries, the 5G module in slot 2 with its SIMs in `J_SIM1`/`J_SIM2` and its pigtails to 5G MAIN and 5G DIV (ANT0 and ANT2), the LimeSDR into `J_LIME` in its bay with its pigtail to SDR, the RockBLOCK on its bracket into `J_RB9704` with its pigtail to IRIDIUM, the GNSS pigtail from `J_GNSS1` to GNSS, the LoRa pigtail from `J_LORA1` to LORA, one module's antenna-kit lead to WIFI 2.4, the CR2032, the four rail leads from A (`J_5V_S1..3`, `J_5V_DEV`), the PoE lead (`J_54V`), the HDMI cable from `J_HDMI` and the camera and QMX leads (`J_CAM`, `J_QMX`) left for the face and the lid, the panel ribbon in `J_PANEL`; the 2x13 `J_AB1` header mates A's at the same case XY as the board comes down. Nyloc on top.
6. Pack into the east pocket (corrected 27 September 2026), cable and SMBus into E.
7. RF: the right-angle plugs sit in their printed clamps on the dock strip and mate blind with the receptacles under A when the stack is lowered. The jumpers from the arrestors' inner jacks run on the routes of `docs/CASE-MARGINS.md` section 3.4 (corrected 27 September 2026), torqued once at the wall side and finger tight at the device side, RG-316 with a 12.5 mm bend radius, tied at both ends.
8. The face (`docs/ASSEMBLY.md` section 2 step 8): press the eight standoffs, the two PA nuts and the sixteen light guides into the plate; the PA module on its thermal pad under the plate with its coax and bias leads to D and its 13.8 V lead to A; the Xenarc on the VESA holes with its block through the cutout and its gasket; the switches, the sounder and the two headset jacks through the plate with their seals, the camera module behind its window, the e-paper taped under the lens; then the backer C onto the standoffs (its LEDs under the light guides, the switch leads to the lands beside each site, the e-paper flex into `J_EPD`, the headset leads to D `J_HS1`/`J_HS2`, the MAIN and PI leads, the ribbon); then the plate onto the frame over Peli's o-ring on its ten 6-32 screws (corrected 27 September 2026, C1). Flood and hose the face in its frame before the stack goes in (appendix 32.34, the same procedure as the previous face).
9. Lid: the QMX tray r2 screwed to its lid plate, which is bonded to the lid's inner face over the right strip, the unit lowered in from above and the retaining frame screwed over it (`docs/ASSEMBLY.md` section 9, sheet 14r2-3), its three leads in the lid harness (USB to B `J_QMX`, 12 V to A `J_HF`, the BNC-to-SMA jumper to the HF arrestor's inside).

Torque table, threadlocker rules and every lead's wire gauge, length and connector are in `docs/ASSEMBLY.md` sections 1 and 4. Never put threadlocker on Nyloc nuts or on the switch nuts.

## 6. Coating and labels

After the bench fit, two thin coats of acrylic conformal coating on A, B, D and E with the masks of `docs/ASSEMBLY.md` section 5 (connector faces, the receptacles and sockets, the spring pins and their targets, SMA and U.FL bodies, the module sites, the test points, the water electrodes on E). The backer's underside is coated after the silicone beads have cured, with `J_PANEL`, `J_EPD`, the lead lands and the standoff rings masked; the plate is bare anodised aluminium. Labels per section 6: the plate nameplate with P/N MSK-FK-1450, S/N, REV A and a data matrix; P/N, S/N, REV silk fields on every board.

## 7. Software

Three Compute Module 5: flash each eMMC with `rpiboot` through B's `J_FLASH` with the `J_RPIBOOT` jumper on the slot being flashed (the B schematic names the strap per slot), Raspberry Pi OS with the carrier's overlays, then k3s across the three (one server, two agents, replicated storage on the NVMe drives) and the HAL (MESHSAT-801) that shares the USB devices cluster-wide. The kit has no radio on a module GPIO except the LoRa module on slot 3's SPI header (`meshtasticd` on `spidev0.1` with BUSY, DIO1 and reset on GPIO 23, 24 and 26): the LG290P, the two E72, the panel controller, the sensor controller, D (a USB audio and control set), the RockBLOCK, the LimeSDR, the QMX and the camera are USB devices on the per-slot hubs; the 5G module's data runs on slot 2's PCIe lane and its management link is USB, and the two WiFi link cards are PCIe cards on slots 1 and 3 (corrected 27 September 2026). Ethernet ties the three modules through the KSZ9897 switch to the wall RJ45. The Xenarc is an HDMI monitor with USB touch behind the three-input display switch that the panel controller selects; the kiosk runs on whichever module owns the display (`docs/PANEL.md` section 5).

- Panel: `docs/PANEL.md` is the contract of the panel controller firmware (MESHSAT-837) and the bridge protocol over USB. Corrected 27 September 2026: until it lands, MAIN PWR and the EMCON gates act in hardware, the indicator rail `LED_RAIL` stays dark, and the TX lamp with it, because C's high-side switch feeds that rail only while the firmware drives `PANEL_PWM` (`docs/PANEL.md` section 3, GPIO 8; `docs/feasibility/EMCON.md` section 0), no compute module runs (the slot enables stay low), and ZEROIZE does nothing, because the erase is the panel controller's firmware and provisioning behind a hardware toggle input (owner ruling D-03; `docs/PANEL.md` sections 6 and 7).
- Sensors: the sensor controller on E (MESHSAT-838) reports the climate, seal, water, gas, motion, lightning, Geiger and outside-pod readings over USB; the alarm rules are the bridge's.
- Power: the charger, the rail monitors and the rail enables are on the kit I2C bus mastered by the panel controller; the bridge reads them through it (SHORE, CHARGING, the battery bar, the per-slot currents) and asks it for the shore inhibit and the slot power cycles.
- The issue list of the software of this generation: MESHSAT-835 to 848 (`docs/V2-SPEC.md` section 7).

## 8. Bring-up checks

`docs/TEST-PLAN.md` is the qualification plan; the first-power checks from `docs/ASSEMBLY.md` section 8: the dock strip gives its 20 V bus with 9, 12, 24 and 36 V in, survives reverse polarity for 10 s and blows its fuse on a bolted short; each slot rail comes up to 5.1 V under 3 A; the lamp test lights all seventeen controller-lit indicators (corrected 27 September 2026: not `D22`, the hardware EMCON lamp, which setting EMCON tests; `docs/PANEL.md` section 9), BLACKOUT kills the rail, the EMCON cover closed keeps the SA868 and the PA in receive while the bridge asserts PTT; the shore inhibit drops and restores the front end and the kit keeps running from the pack (record the current, it sets the survival time); at full load measure the current on the block's return pins against the pin rating; the PA flange temperature after a key-down at 30 W into a load (corrected 27 September 2026: a PA key-down is bounded at 60 s, PROVISIONAL, session choice SC-10, and on the design record's own figure the flange passes the maker's 90 C reliability figure within that time from a +50 C plate, so the flange is watched with a thermocouple, `docs/feasibility/POWER-THERMAL.md` finding PWR-F15). Then the V1 checks (`../v1/BUILD.md` section 8) for the radios, the modem, the display and the demo.

Removal for maintenance (`docs/ASSEMBLY.md` section 7): lid, the ten plate screws, the ribbon, the headset and PA leads, the face out, then lift the A + D + B stack straight up. Nothing has to be unscrewed at the radio side: the RF joints and the power contacts part as the stack rises, and the rods through the dock strip line them up again on refit. Before the lift the kit is off, the pack's XT60 unplugged and shore removed, and an insulating cap covers the dock block E5 while the stack is out (corrected 27 September 2026, owner ruling D-14).

## 9. Known gaps of this generation

- Nothing here has been built and no board has been fabricated. Report what does not fit on MESHSAT-830.
- Corrected 27 September 2026: the foundations beneath the boards are incomplete and no board is ready for layout (`docs/CURRENT-EVIDENCE.md`); the circuit corrections of 26 September 2026 are in the schematics only, and every deliverable folder predates them.
- The sealed face (the plate with C under it) is a construction, not a test result: the flood, hose, rain and dust procedure of appendix 32.34 has not been run on any face; the whole-kit MIL-STD-810 and 461 programme of `docs/TEST-PLAN.md` has not started.
- Corrected 27 September 2026: the pack is one shrink-wrapped 4S3P block in the east pocket by owner ruling D-06; its board P is generated, the D-15 second level is in its schematic only, the block's welding and the gauge's golden image are bench work after the D-09 review, and no second pack has a location (D-01 defers it).
- Part picks owed: the toggle safety covers, the U-174/U jacks' drawing, the camera module, the sealed RJ45 and USB-C wall parts, the fans, the tablet, the 2 m antenna (the laptop research list of appendix 32.49); the NVMe drives' grade and the two bought parts not rated to the envelope's -20 C (the WiFi link cards, from 0 C or -10 C as the maker's two documents disagree, and the LimeSDR, from 0 C; `docs/feasibility/POWER-THERMAL.md` section 9.4).
- The QMX in the lid tray is a session decision under the owner's requirement for an HF unit inside the case (appendix 32.60 item 5, veto open); the tablet bracket is not drawn.
- The PA's thermal path (the flange on the plate) is an estimate until a module is keyed on a plate; the 30 W stage, the T/R relay and the LPF of D have not been measured.
- The three-module fabric (PCIe switches, USB 3 hubs, the HDMI and Ethernet switches) is generated from the makers' reference designs and has not been powered; the module's boot from its eMMC through this carrier, the display switch and the HAL sharing are bench items.

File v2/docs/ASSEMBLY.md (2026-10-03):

# MeshSat Field Kit carrier set: assembly, fasteners, coatings, removal (Rev A, MESHSAT-830)

Companion to `MESHSAT-709-geometry-appendix.md` (sections 32.49 to 32.61) and `../BUILD.md`. Boards: PCB-A POWER + I/O (**A22**), PCB-B COMPUTE (**B16**), PCB-C PANEL BACKER (**C7**, the ring under the aluminium face plate), PCB-D VHF APRS (**D8**, the mezzanine on A22), PCB-E1 DOCK STRIP (**E6**, with the sensor controller on it), PCB-E5 DOCK BLOCK (**E5**). Nothing here has been built; this is how the first set is meant to go together. The previous generation's page (the twelve-cell battery module, the previous display, the single Compute Module) is in the git history of this file.

The set of 7 September 2026: three Compute Module 5 slots on B16 with a PCIe switch, a USB 3 hub and an NVMe drive each, the radios as USB devices, an Ethernet switch to a sealed wall port, the Xenarc 709GNK monitor set into the face plate with its glass level with the aluminium, the Pervasive Displays e-paper under a lens, the RP2040 panel controller on C7, the SA868 exciter and the RA30H1317M1 30 W amplifier (the module bolted under the plate) on D8, a built 4S smart pack in the pocket at the east wall (appendix 32.62), the 9 to 36 V front end and the solar tracker on E6, eleven blind-mate RF paths through the dock, and the QMX HF unit in a tray on the lid.

> **Corrections of 26 September 2026 (MESHSAT-1357), each marked where it is made.** Read against the generators
> and the committed boards at `82dd1e4d`; nothing has been built, so each is a correction to the design record,
> not to a kit. (1) D8 sits on 6 mm standoffs, not 22.6 mm ones: 22.6 is the Z of D8's underside. (2) A22's
> `J_AB2` header stands under D8 and is expected to collide with it on those standoffs: an OPEN design finding
> (INFERRED from the header's class height, section 1). (3) The A22 to B16 bay spacers are about 31.3 mm, not
> 38 mm, since B16 dropped to its current height on 9 September (INFERRED until the stack is drawn, section 1).
> (4) The RockBLOCK bracket sits on four M4 holes, not M2.5. (5) No 4S pack of the sizes section 3 promised is
> expected to fit the east pocket beside the pack board, no rigid enclosure is expected to fit at all, and no
> pack is expected to fit the west pocket (INFERRED from the committed board heights, section 3; the case side at the worst of Peli's figures, `CASE-MARGINS.md`); the owner has ruled
> the pack to fit that finding (D-06). (6) The pack's SMBus lead had no single connector: the two ends were
> different families with different pin orders (superseded by `faf8c981`, see (12)). (7) The charger has no thermistor input; the pack's gauge holds
> charging off on its own. (8) The stack is never lifted live: the dock-lift procedure and the insulating cap
> over E5 are the owner's ruling (D-14, section 7). (9) The wall data path moves to the sealed Glenair and the
> USB-C outlet becomes power only (D-12, section 4); the generators did not do that yet (superseded by `458b2873`, see (12)). (10) The 5G antenna
> jacks are ruled at three (D-07; its case condition is answered by `CASE-MARGINS.md` section 3.4 after the owner reversed D-08, the board E clamp fit remains), which makes twelve bulkheads; the
> eleven RF paths this document counts are the generated set and change with that board work. (11) Later on 26 September 2026 (appendix 32.367): the owner reversed D-08 at about 09:30 CEST, so no case measurement and no mock-up are asked of him, and every fit that waited on them is designed against the worst of Peli's own figures (`CASE-MARGINS.md`), with the margins that rest on a tolerance no source states OPEN until a targeted unpowered mock-up at the build stage (that timing is replaced by item (13) of 27 September 2026); the design targets the current moulding of Peli's drawing 1451-931 of 15 January 2025 (D-08a). Items (5) and (10) and section 3 are corrected to match.
> (12) Later on 26 September 2026 (open item S-07 of the requirements registry), read against the generators and the
> committed netlists at `45bde541`, which carry the circuit corrections of `faf8c981`, `458b2873` and `d90f30e4`: the
> SMBus lead is one JST-XH 1x4 at both ends in board P's order; the wall data path leaves A22 at `J_USBW` for the
> Glenair and the USB-C outlet carries power and CC only, with an ESD array on its CC pins; the heater mat gets a
> regulated 12 V; the second WiFi link card on slot 3 and the antenna changeover the two cards share are in the build
> and lead lists; the pack lead is board P's own, not the withdrawn BB-2590/U cable; board P carries the second level
> and chemical fuse of D-15, armed at commissioning; the charger's strap selects 4S; a lid and tamper reed switch is on
> E6. Section 2 steps 1, 6 and 7, section 4 (its rows and the dock paragraph), section 8 steps 4 and 12 and section 9
> are corrected to match, each where it is made. Nothing of it is laid out or built.
> (13) 27 September 2026 (MESHSAT-1357, pre-PCB layer 7): the case set `v2/release/case-2026-09-27/` (STEP, DXF, dimensioned
> drawings, 1:1 templates, generated from `v2/ecad/tools/panel1450.py`) implements the session's choices C1 to C6 (SC-07,
> `CASE-MARGINS.md` section 4). The rows of sections 1 to 4, 6, 7 and 9 that named the face plate on M3 from below with a PORON
> ring, the connector plate between ribs, the Amphenol couplers at Z 88, the stack's old heights, the QMX tray at X 103.5, the lid
> space and the pack's pocket are corrected to it, each marked where it is made; the QMX tray's part and place are sheet 14 and
> `lid-tray-qmx/` of that set (added by the layer 7 fixer c7 the same day). The targeted mock-up's checks of the rows that can move
> a board (the YES rows of `CASE-FIT-UNCERTAINTIES.md` section 2) are **required before the layout entry of boards A, B, E and P**,
> and that layout entry is BLOCKED on the owner's purchase decision (D-09; FEA-007; `CASE-MARGINS.md` section 7 as revised on 27
> September 2026, `CASE-FIT-UNCERTAINTIES.md` section 7); boards C, D and E5 are not held by it, and the other checks run at the
> build. This replaces the build-stage timing of item (11) and section 3, and the seventh revision's recommendation (before the
> outlines of A, B, C, E and P freeze). Still owed, and listed with the check each waits on in `CASE-FIT-UNCERTAINTIES.md`: the jumpers' right-angle
> plug (M17g and M17x fail with the plug as laid out), the pack's hold-down (S-27), the rod stack's retention (W4-F7), the dock and
> blind-mate tolerance stack, the fans and the floor plan, and the QMX tray's fit to the unit (its fastener row; answered by the r2 set on 27 September 2026, whose verification is S-96 and whose leads' crossing of the face is S-95). Nothing of it is
> made, bought or fitted.

## 1. Fasteners

| Joint | Fastener | Torque | Locking |
|---|---|---|---|
| Rod stack, 4 x | M3 stainless threaded rod, floor to the top nut above B16; spacer tubes on the dock strip that set the 13.4 mm blind-mate gap under A22; bay spacers between A22 and B16 of about 31.3 mm (corrected 26 September 2026: this read 38 mm with B16's top copper at 56 mm, the figures before 9 September). **Corrected 27 September 2026 (MESHSAT-1357, the case set C1 to C6):** the stack is drawn from the boards (`panel1450.py` STACK; the Z-stack sheet 5 of `v2/release/case-2026-09-27/`): the dock strip's VHB 5952 pads 1.1, E6 1.6, the gap spacer 13.4, A22 1.6, the bay spacer 31.3, B16 1.6, so A22's top is at Z 17.7, B16's underside at Z 49.0 and its top copper at Z 50.6; the gap and bay spacers are still unnamed parts (TBD, `CASE-MARGINS.md` section 6), and the north rods have no foot (W4-F7, the retention is not designed) | 0.5 N m | Nyloc nuts top and bottom, no threadlocker on Nyloc |
| Face plate to frame, 10 x (Peli 1450PF) | **Corrected 27 September 2026 (MESHSAT-1357, the case set C1 to C6):** 10 x 6-32 UNC x 1/2 in A2 pan head (ASME B18.6.3 class, 6.86 across the head at most) from above, by hand, through the plate's 4.6 mm holes into Peli's brass inserts at the frame STEP's bores (X +-179.07 at Y +-75.95; X 0 and +-139.45 at Y +-121.16); the 377.2 x 263.0 plate lies on the frame's top face and covers Peli's o-ring in the channel between the frame and the case wall (Peli's mounting instructions, steps 2 to 4); no PORON ring (C1, `v2/release/case-2026-09-27/face-plate/`). Until 27 September 2026: M3 x 10 from below with a PORON 4701-30 ring | hand tight, no pressure (Peli's instruction); a torque is TBD from Peli | none (Peli's inserts); T3 dry-fits it |
| Setting legs to the frame, 4 x | **Corrected 27 September 2026 (MESHSAT-1357, the case set C1 to C6):** one 6.0 mm 6061-T6 leg under each corner of the frame's ring (C6, `v2/release/case-2026-09-27/frame-legs/`), bonded by a 3M VHB 5952 pad in the 0.9 mm pocket of its pad top so the aluminium rim, not the tape, meets the ring; placed with the frame face down on the bench by the printed locator that drops into each window corner; the feet stand bare on Peli's floor, pad top 94.13 +-0.10 above the foot | pressed as 3M's VHB guidance asks (TBD from its sheet) | the bond (T8 tests VHB on the frame's polymer, which Peli does not state) |
| 1450PF frame to the case, 4 x | **Corrected 27 September 2026 (MESHSAT-1357, the case set C1 to C6):** Peli's four self-tapping screws through the skirt, as Peli instructs, after the frame on its legs is centred by two pairs of printed wedges (0 to 2.0 over 40) pushed to equal depth marks at the middles of opposite walls; the wedges come out, then Peli's o-ring goes into the channel | Peli's | none |
| Backer C7 to the plate, 8 x | M3 x 6 A2 into the eight PEM SO-M3-10 self-clinching standoffs pressed into the plate from below (4.2 mm holes; `panel1450.py` STANDOFFS), through the backer's GND rings H1 to H8, which bond the backer to the plate | 0.4 N m | Loctite 243 |
| PA module to the plate, 2 x | Mitsubishi RA30H1317M1 flange under the plate at `PA_MOUNT` (flange holes 60 mm apart, 3.26 mm), M3 x 8 into two PEM S-M3 nuts pressed into the plate's underside, a 1.0 mm thermal pad the size of the flange between module and plate; the plate is the heat spreader (appendix 32.56) | 0.6 N m in two steps | Loctite 243 |
| Xenarc 709GNK in the plate, 4 x | The monitor drops into the plate's 205.75 x 140.09 R15 window from above until its **glass surface is level with the plate's top face** (owner ruling 9 September 2026, appendix 32.85 and 14.6): its 10.66 mm bezel flange fills the plate's 3 mm and its 18.00 mm rear shell hangs into the void. A closed-cell foam gasket seals the flange to the window land all round; a steel rear frame under the plate, M4 x 8 at the four `XENARC["frame_holes"]`, pulls the monitor up against it and carries the 1.2 kg (the monitor's own VESA 50 inserts take M4 x 6 mm maximum, so the frame is the load path, not the plate) | 1.0 N m | Loctite 243 |
| Light guides, 17 x | Mentor 1282.5004 (IP68, 2.5 mm shaft, 3.2 mm spherical head, 7.5 mm long) pressed from the face into the 2.6 H7 reamed holes over D1 to D16 and D22; the LEDs on the backer stand 5.3 mm high, 0.2 mm under the guide tips. D22 is the hardware EMCON lamp that board C's round 8 of MESHSAT-1357 (26 September 2026) draws beside `SW_EMCON` (SD-EMC-6); its hole is not yet in the plate (`panel1450.py`) and its position is placed at board C's next layout | press fit | none |
| Connector plate to the back wall, 6 x | **Corrected 27 September 2026 (MESHSAT-1357, the case set C1 to C6):** M4 x 25 A2 at X +-51.1, Z 24.2, 50.1 and 76.0 through the back wall between the hinge fairings (the 114.0 x 68.3 x 5.0 plate centred at X 0, Z 18.3 to 86.6, C3; `v2/release/case-2026-09-27/connector-plate/` and the back-wall template, sheet 1 of `templates/case-templates-1to1.pdf`), a bonded sealing washer 10 across under each outside head, a plain washer and a Nyloc inside, a 2 mm closed-cell gasket of the plate's outline between plate and wall. Until 27 September 2026: M4 x 16 between inner ribs at X -95 and -18 that Peli's files do not show | 1.2 N m (TBD from the sealing washer's maker) | Nyloc |
| RF entry plates to the end walls, 2 x 8 | **Corrected 27 September 2026 (MESHSAT-1357, the case set C1 to C6):** M4 x 12 A2 ISO 7380 button heads from inside through the wall's 5.0 mm holes into threads tapped through the 6.0 mm plate at Y +-45 and +-100, Z 40.65 and 77.35, each on a rubber-faced sealing washer 10 x 1.5 (face 8.0 across or more) over its hole; a 2.0 mm closed-cell gasket of the plate's outline (220.2 x 48.9, Y +-110.1, Z 34.55 to 83.45) between plate and wall (C4, `v2/release/case-2026-09-27/rf-entry-plates/`, templates sheets 2 and 3) | none stated (TBD from the sealing washer's maker, `CASE-MARGINS.md` section 6) | none |
| Arrestors on the RF entry plates, 5 east + 7 west | **Corrected 27 September 2026 (MESHSAT-1357, the case set C1 to C6):** PolyPhaser GTH-SFF-AL through the plate's 16.3 mm holes, its own O-ring on the plate's machined outer face, its lock washer and nut on the floor of the 26.0 x 1.5 spot-face in the plate's back, cap up and ground lug down; tightened on the bench before the plate goes on the wall (a 30 mm socket clears the next nut) | the maker's (not on its sheet, TBD) | the lock washer |
| D8 on A22, 4 x | M3 x 6 into four **M3 x 6 mm** standoffs at A22's mezzanine site (5, +-35) and (95, +-35) (`gen_pcb_a.py` MEZZ_RECT), which puts D8's underside at Z 22.6, 6.0 mm above A22's top at 16.6 (appendix 32.85, `scene.py:275`; corrected 26 September 2026, this row gave 22.6 mm as the standoff length). **OPEN design finding, 26 September 2026:** A22's `J_AB2`, the vertical 2x5 wall-port ribbon header added on 12 September (`gen_pcb_a3.py:74`, at (95, -11) inside MEZZ_RECT 0 to 100 by -40 to 40), stands under D8. Its body is about 9.1 mm tall (INFERRED: it has no picked part, and 9.1 mm is its DIN 41651 class) in a 6.0 mm gap, so D8 is not expected to seat (INFERRED), and no single standoff height is expected to clear both `J_AB2` below and B16 above (INFERRED from the 31.3 mm bay). No gate checks heights under the mezzanine. Either `J_AB2` moves out of the mezzanine rectangle or D8's height is re-derived from both sides | 0.5 N m | Loctite 243 |
| Compute Modules on B16, 3 x 4 | M2.5 x 4.0 female-female standoffs on each module's 33 x 48 pattern (the height of the 10164227-1004 receptacle stack), M2.5 x 5 from below, M2.5 x 4 from above; the CM5 Cooler clips on each module, its fan lead in `J_FAN1..3` | 0.2 N m | Loctite 243 on the standoff thread only |
| M.2 cards on B16, 6 x | M2.5 x 4.0 standoff at the far end of each socket (`J_M2C1` E-key 2230, `J_M2C2` B-key 3052, `J_M2C3` M-key 2242 spare, `J_M2N1..3` M-key 2242 NVMe), M2.5 x 4 screw | 0.2 N m | none |
| RockBLOCK 9704 on B16 | the Ground Control bracket on four **M4** standoffs, 8 mm, over B16's 4.3 mm holes H17 to H20 on a 32 x 32 pattern (`gen_pcb_b.py:187`, "M4, GC 9704 bracket"; corrected 26 September 2026, this row said M2.5), the 2x8 IDC lead to `J_RB9704`. The fasteners below B16 reach into the east pack pocket and their type and drop are still owed | TBD for M4 (0.2 N m was the M2.5 figure) | none |
| LimeSDR Mini in its bay | plugged into the USB 3 A receptacle `J_LIME`; a cable tie base beside the bay and one tie over the board keep it seated | | tie |
| E-paper under the plate | Pervasive Displays E2370KS0C1 face-up under the plate, glass up in the 94.19 x 53.6 window, its side lands taped to the plate's underside with 3M VHB 5915; in the plate's 1.0 mm top pocket a **1.0 mm** UV-grade polycarbonate lens 107.19 x 66.6 on a 6 mm die-cut frame of 0.05 mm acrylic transfer tape (3M 467MP or 9495LE), 3M Primer 94 on the lens's bonded face, so the lens ends **0.05 mm proud** and meets the ruling of 14.6 that every display surface is level with the face; foam tape anywhere here breaks that limit; the 24-way flex leaves the left short edge into `J_EPD` on the backer's top strip; no screws | | tape |
| Panel switches (in the plate, their bodies through the backer's slots and holes) | supplied nuts; SW_MAIN, SW_PI, SW_TEST on a die-cut 1.0 mm Silex GP60 silicone washer under the bezel; SW_LIGHT (NKK D3 bushing) with its O-ring (spare AT516) under the nut on the face and the AT428H boot, its D flat east; SW_SOS, SW_EMCON, SW_ZERO with the APEM K seal keyed into the notch toward the operator and the hinged safety covers on SOS and ZEROIZE (cover part owed); flying leads soldered to the backer's lands beside each site, then beaded | hand tight + 1/8 turn | none |
| Headset jacks, 2 x | U-174/U panel jacks (Amphenol Nexus class, drawing owed) through the plate's holes at `HEADSETS`, bushing nut below the backer's 17 mm holes, sealing washer on the face; five-lead pigtail to D8 `J_HS1`/`J_HS2` | hand tight | none |
| Camera module | the USB camera board (about 25 x 25 mm, part owed) on two M2 standoffs behind the plate's 8 mm sealed window at `CAMERA` (`CAM_H1`/`CAM_H2` on the backer), the window glazed from the outside with a 1.0 mm PC disc on VHB 5915; its USB lead to B16 `J_CAM` | 0.15 N m | none |
| Light sensor window | the VEML7700 on the backer under its own Mentor light guide in the plate at `LIGHT_SENSOR` | press fit | none |
| Sounder BZ1 | Floyd Bell MC-09-530-Q through the plate's 28.6 mm hole with the 61663 bezel gasket on the face, nut below the plate, two leads to the lands | hand tight | none |
| QMX tray on the lid (r2), 10 x and 6 x | **Replaced 27 September 2026 (MESHSAT-1357, S-63, SC-TR-01): the r2 set** `v2/release/case-2026-09-27/lid-tray-qmx-r2/` (sheets 14r2-1 to 14r2-3; the r1 tray of `lid-tray-qmx/` and sheet 14 are superseded and not printed): a 2.0 mm 5052-H32 lid plate (`lid-plate-qmx-r2.dxf`, ten M3 tapped through) bonded to the lid's unribbed inner face with 3M DP8005 at case X 83.2 to 171.0, Y -45.9 to 65.9 (its east edge where C5 put r1's, M19 unchanged); the tray, printed in Prusament PC Blend (100 percent infill, 0.20 mm layers), on it with ten M3 x 5 countersunk hex socket (ISO 10642 class) A2; two Rogers PORON 4701-30 pads (3.18 mm, 24 x 20) in the floor windows; the unit, without its optional rubber feet and with its knobs on, top face out, its knob edge west and its right panel (RF, PTT, USB) toward the hinge, LOWERED INTO THE POCKET FROM ABOVE; the retaining frame (PC Blend, flat, 3.0) laid over it on the wall tops and screwed with six M3 x 10 button head (ISO 7380-1 class) A2 into six M3 square nuts (DIN 562 class) in the posts' slots, which compresses the pads by 1.08. Both end panels stay open: every jack takes its plug (`lid-tray-qmx-r2-check.out` section A) | 0.25 N m on all sixteen (INFERRED; the r1 row's 0.4 N m would load 1.4 mm of thread in 5052 to 67 percent of what it strips at) | a threadlocker whose maker states it compatible with polycarbonate (the pick is TBD; r1 named Loctite 243 for a PETG tray) |
| Dock strip to floor | 4 x 3M VHB 5952 pads 20 x 20 at the corners, floor degreased with IPA | | |
| Pack to floor | the pack on four VHB 5952 pads in the east pocket (from board A's edge at X +120 to Peli's floor fillet and east wall, under B16's overhang, centred in Y so that each end keeps 3.65 mm to the frame's setting legs, 1.77 at the worst, `CASE-MARGINS.md` M4a to M5), the RS PRO 245-556 heater mat stuck to the floor under it. **Corrected 26 September 2026:** the printed enclosure of `v2/cad/pack_4s.py` (56 x 236 x 46) is not expected to sit in this pocket under B16: it meets B16's underside `J_AB2` header and U.FL cluster, and no rigid enclosure is expected to hold a 4S block with the pack board in this pocket (INFERRED from the committed board heights, section 3). The owner's pack ruling (D-06) is a shrink-wrapped 4S3P block here; how it is held against the drop and vibration tests (`TEST-PLAN.md` E1, E2) has not been designed or assessed | | |
| Blade fuses | 25 A mini blade in A22 `F1` (the pack node), 25 A in E6 `F3` (pack), 10 A in E6 `F1` (vehicle input) and `F2` (solar), Keystone 3568 holders | push fit, seated flush | none; check seating after any transport |
| Dock block E5 | four M3 x 6 standoffs above the strip, face at 7.4 mm (**Corrected 27 September 2026 (MESHSAT-1357, the case set C1 to C6):** a 6.0 standoff under the 1.6 block puts its face at 7.6, not 7.4; the dock and blind-mate tolerance stack names the standoff, `CASE-FIT-UNCERTAINTIES.md` section 3, row DOCK) | 0.4 N m | Loctite 243 |

Threadlocker: Loctite 243 (medium, oil tolerant) on every machine screw into metal; never on Nyloc nuts, never on the plastic-bodied switch nuts.

## 2. Build order

0. **Corrected 27 September 2026 (MESHSAT-1357, the case set C1 to C6):** the case first. Drill and saw the wall holes from the 1:1 templates (`v2/release/case-2026-09-27/templates/`: the back wall's 29, 22, 18 and 8 mm holes and six 4.5 mm; each end wall's 27 mm hole-saw holes at the arrestor sites and eight 5.0 mm), deburred; the connector plate with its six items on its gasket (section 1); the arrestors tightened on their RF entry plates on the bench, then each plate on its gasket on its end wall. Bond the four setting legs under the frame's ring with the locators (frame face down on the bench), lower the frame on its legs into the case, centre it with the wedges, drive Peli's four screws, take the wedges out and fit Peli's o-ring in its channel. The frame and its legs stay in the case from here on; the dock strip, the stack and the pack go in through the frame's window (349.65 x 233.83), and the face plate goes on last (step 9).
1. Dock strip E6: solder the entry leads (vehicle and shore pair to `J_DCIN`, solar pair to `J_SOLAR`, VH crimps), the pack cable's XT60 counterpart at `J_BATT` and the SMBus socket `J_SMB` (JST-XH 1x4), the lid and tamper reed's lead into `J_TAMP`, the sensor headers (`J_DCF`, `J_GEIGER`, `J_LTG`, `J_POD`), the two mixer fans (`J_FAN1`, `J_FAN2`), the water electrode leads; fit the three fuse holders with their blades, and check the 20 V bus at the block lands with 9 V and 36 V in. The front end, the tracker and the sensor controller are assembled parts.
2. Dock block E5 on its four M3 x 6 standoffs above the strip. Solder the twelve signal wires and the 12 AWG pair from the strip into the block's plated lands from below; the block's underside legend names every land. Check each wire end to end before the stack goes on, because the lands are covered once A22 is down.
3. Rods: four M3 rods through the floor holes of the strip, then the spacers that set the 13.4 mm gap on all four rods, so A22's spring pins land on the block with the pins compressed about 1 mm.
4. A22 with the Preci-Dip 813-S1-012-10-016101 connector and the seventeen Mill-Max 0858 class power pins (nine for the pack, `J_CP1` to `J_CP4`, `J_CN1` to `J_CN4` and `J_PRE1`, and since EQ-16 eight for the input, `J_VR1` to `J_VR4` and `J_VN1` to `J_VN4`) soldered in from the underside (tails on the top face), the eleven Radiall receptacles fitted, and the blade fuse in before anything is energised. Lower it onto the rods and check continuity from the block's wire lands up to the board.
5. D8 onto A22's four 6 mm standoffs (D8's underside at Z 22.6; corrected 26 September 2026, and blocked by the open `J_AB2` finding of section 1): the 2x8 harness ribbon `J_MEZZ1` to `J_HARN1`, the 5 V lead `J_MEZZ_PWR1` to `J_PWR1`, the antenna pigtail from `J_ANT` to A22's VHF jack `J_RF1`; the PA drive coax (`J_PAIN`), the PA output coax (`J_PAOUT`), the gate bias lead (`J_VGG`) and A22's 13.8 V lead (`J_PA`) coiled and tied for the plate.
6. The bay spacers (about 31.3 mm, section 1; corrected 26 September 2026 from 38 mm), B16: the three Compute Modules pressed onto their receptacle pairs and screwed to the standoffs, the coolers clipped on with their fan leads in `J_FAN1..3`, the NVMe drives in `J_M2N1..3`, the two WiFi link cards in `J_M2C1` (slot 1) and `J_M2C3` (slot 3), each with its two MHF4 pigtails to B16's antenna changeover (`J_W1A`, `J_W1B` and `J_W3A`, `J_W3B`), the changeover's two outputs (`J_WOA`, `J_WOB`) by pigtail to A22's P2P A and P2P B jacks, the 5G module in `J_M2C2` (slot 2) with its SIMs in `J_SIM1`/`J_SIM2` and its pigtails from its ANT0 and ANT2 receptacles to the 5G MAIN and 5G DIV jacks (ANT3, the third jack of D-07, waits on A22's site; corrected 26 September 2026, S-07: this step named one card and pigtails straight to the wall), the LimeSDR into `J_LIME` with its pigtail to SDR, the RockBLOCK on its bracket into `J_RB9704` with its pigtail to IRIDIUM, the GNSS pigtail from `J_GNSS1` to A22 `J_RF4`, the LoRa pigtail from `J_LORA1` to `J_RF11`, one module's antenna-kit lead to `J_RF3`, the CR2032, the four rail leads from A22 into `J_5V_S1..3` and `J_5V_DEV`, the PoE lead into `J_54V`, the 26-way ribbon between A22's and B16's `J_AB1` (the two headers sit at the same case XY, one on A22's top and one on B16's underside), the HDMI cable in `J_HDMI` and the camera and QMX leads in `J_CAM` and `J_QMX` left for the face and the lid, the panel ribbon in `J_PANEL`. Nyloc on top.
7. Pack into the east pocket (its hold-down waits on the redesign of `v2/cad/pack_4s.py`, section 3), the pack lead's XT60 (board P's own two 12 AWG leads from `W_P` and `W_N`, `gen_sch_p.py:347-348`) into E6 `J_BATT`, the SMBus lead's XH housing into `J_SMB` (a straight four-way XH lead, pin n to pin n, section 4). Board P's chemical fuse stays disarmed (its jumper `JP1` open) until commissioning, section 8 step 12. **Corrected 26 September 2026 (S-07):** this step named the BTA-70762-2 cable of the withdrawn BB-2590/U, which `J_BATT`'s value text in `gen_sch_e.py:193` still carries at `45bde541` (a stale label for board E's writer).
8. RF: the right-angle plugs sit in the cavities of the printed float clamp bar on the strip (one bar for every site since 26 September 2026, A09 and R4E-07; twelve cavities, the twelfth for D-07's third 5G jack at X +46, which takes a plug once board A carries its receptacle) and mate with the receptacles under A22 as the stack comes down. The wall pigtails run from the clamps to the end-wall couplers, torqued once at the wall side and finger tight at the device side. **Corrected 27 September 2026 (MESHSAT-1357, the case set C1 to C6):** the jumpers (RG-316, each cut to its route of `CASE-MARGINS.md` section 3.4 plus 20 mm, 252 to 432 mm) run from the clamps to the arrestors' inner jacks on the RF entry plates, a right-angle SMA male crimp plug on each: on the east wall each plug turned 30 degrees below the wall's direction toward its bundle's end (5G MAIN, 5G DIV, 5G ANT3 and IRIDIUM in a front bundle, LORA in a back one, over the pack's outer strip, inboard of the legs' columns and down beyond the legs), on the west wall each cable straight down; every bend at R 12.5 or more. The plug is not picked, and with the plug as laid out two east rows fail (M17g, M17x): the pick decides board B's east edge (`CASE-FIT-UNCERTAINTIES.md` section 2), and T10 lays the real jumpers. The ANT3 path waits on its site on A22 and a clamp at X +46 on E6 (D-07).
9. The face (appendix 32.56, 32.60): press the eight PEM standoffs, the two PA nuts and the sixteen light guides into the plate; the PA module on its thermal pad under the plate with its two coax leads and the bias lead to D8 and the 13.8 V lead to A22; the Xenarc lowered into its window from above onto its gasket, then the rear frame drawn up under the plate until the glass is level with the aluminium; the switches, the sounder and the two headset jacks through the plate with their seals, nuts from below; the camera on its standoffs behind the window; the e-paper taped under its window with its lens on the tape frame in the top pocket; then the backer onto the standoffs (its LEDs under the light guides, 8 x M3 x 6), the e-paper flex into `J_EPD`, the switch and sounder leads soldered to the lands beside each site, a bead of DOWSIL 3145 over the LED joints and every lead land, cured; the backer's underside coated (section 5); the MAIN lead to A22 `J_MAINSW` and the PI button leads to `J_PIJ2`'s lands, beaded; the headset pigtails to D8; the HDMI, USB touch and 12 V leads of the monitor below the plate to B16 `J_HDMI`, D8 `J_USB3` (the touch lead through its USB A to PH 1x4 adapter, section 4; the session's choice SC-HF-06 of 27 September 2026, `HW-FW-CONTRACT.md` section 8) and A22 `J_MON`; the ribbon into `J_PANEL`; **Corrected 27 September 2026 (MESHSAT-1357, the case set C1 to C6):** the plate onto the frame's top face over Peli's o-ring, ten 6-32 UNC x 1/2 in from above into Peli's inserts, by hand (C1); no PORON ring and no screw from below. The face's water tests run on the mock-up case with nothing inside that a leak can harm (T7: `TEST-PLAN.md` E6 and E7), not on a frame out of its case as this step said before C1.
10. Lid (**r2, 27 September 2026**): the lid plate bonded with DP8005 (clamped 2 h), the tray screwed to it, the pads laid in, a square nut in each of the six slots, the unit lowered in from above with the lid held level, and the frame screwed over it (the QMX tray row above; sheet 14r2-3 note 1); its USB-C lead to B16 `J_QMX`, its 12 V lead to A22 `J_HF` and its BNC-to-SMA jumper to A22's HF jack `J_RF2`, each tied within 60 mm of its plug to a tie mount bonded to the lid so that no lead pulls on a jack, the three in one lid harness tied along the hinge side with a service loop (as installed the RG-316 turns at R 12.5 and the DC and USB leads at R 20, so each lead's own least bend radius must be no larger than that; the harness's crossing of the sealed face is not designed yet, S-95, EQ-31). The Paddle, Audio and PTT jacks are the operator's and are unplugged before the lid closes.
11. Lower the lid. Nothing on the face stands more than 0.05 mm proud since the monitor was recessed (9 September 2026), so the whole space between the plate and the lid's inner face is free (**Corrected 27 September 2026 (MESHSAT-1357, the case set C1 to C6):** 47.92 mm nominal from the face top at Z 106.52 to the lid's inner ceiling at Z 154.44, 44.39 at the worst; it read 46.5 before C1); the QMX tray hangs 28 mm from that face and its plan window was sized against the old boxed monitor's east edge, which no longer constrains it (appendix 32.60 item 5, 32.85). **r2 (27 September 2026):** with its lid plate the set's frame stands 32.30 below the ceiling, its six screw heads 33.95, the unit's top face 29.30 and its knob tips 40.90 (knob 11.6, INFERRED). Every face part under the set has its own row in `lid-tray-qmx-r2-check.out` section B, from the deepest solid over it and the part's height from its maker's sheet: the three buttons stand under the frame with heads of 3.50 and 2.50 (C&K ATP19 and ATP16 with their O-rings), 7.96 and 8.96 mm clear at the worst; the knob tips are 3.06 over the flat face and 2.26 over the monitor's window at the worst, 0.35 and -0.45 with every unstated allowance taken twice, so the two knob rows are OPEN until T9; the knobs sit west of the buttons' column.

## 3. The pack

The pack is built for the kit (appendix 32.62; the BB-2590/U of the 6 September ruling is 112 mm tall standing and needs 127 x 112 mm lying, and neither fits beside this board set): a 4S block of sixteen 18650 cells (4S4P, about 200 Wh, about 850 g of cells) or twelve 21700 cells (4S3P), spot-welded on 0.15 x 8 mm nickel strip, with the BMS board P1 (`pcb-p-pack`: the BQ4050 SMBus gauge, protection and balancing, two high-side N-FETs, the 2 mohm shunt, the cell thermistor on TS1), a 25 A mini blade in the board's holder, the printed enclosure with a lid on four M3 corner posts (`v2/cad/pack_4s.py`, `release/revA/case/pack-4s/`: 56 x 236 x 46, the cell block pocket at one end, the board bay on four M3 bosses at the other, a cable notch, two strap slots). It lies in the east pocket beside A22 under B16's overhang (X +120 to +178, Y -120 to +120, Z 1 to 49, the six east-wall couplers well above it) on four VHB pads with the heater mat under it, and connects through an XT60 lead and an SMBus lead of 350 mm along the front wall to E6's `J_BATT` and `J_SMB`. A second pack of the same construction fits the west pocket (58 x 160 x 48) later. Samsung's specification forbids soldering to the cell can: the cells are welded and the leads are soldered to the strip, never to a cell.

**Corrected 27 September 2026 (MESHSAT-1357, the case set C1 to C6):** the pocket is bounded by board A's east edge at X 120 and by Peli's R 15.88 floor fillet and east wall (X 178 is not a Peli surface); B16's underside is at Z 49.0 with the dock strip's VHB pads under the stack (it read 47.9); the block's west face is at X 122.0 and the group (block, board P, 2.0 between) is centred in Y between the east setting legs (`panel1450.py` PACK_BLOCK, PACK_WEST_X, PACK_GROUP_LEN; sheet 6 of `v2/release/case-2026-09-27/`); the east-wall bulkheads are the arrestors at Z 59 on the RF entry plate, whose bottom screw heads keep 3.18 mm to the block's east face at the worst (M4c). The hold-down is not designed (S-27): M4a and M5 wait on it, and `v2/cad/pack_4s.py` is superseded.

**Corrected 26 September 2026: the paragraph above does not fit the board set as it stands.** Measured on the committed B21 board's underside heights (B16's underside is now at Z 47.9, not the 54.4 behind "Z 1 to 49"), with the pack board P, the heater mat and the VHB pads in the same pocket, and every fit INFERRED from the committed board heights, the case side at the worst of Peli's own figures (`CASE-MARGINS.md`):

| pack | east pocket (58 x 240) | west pocket (58 x 160) |
|---|---|---|
| 4S4P 18650, about 193 Wh | does not fit in any packaging tried with board P beside it (the shortest block with the board at its end is about 32 mm too long) | does not fit |
| 4S3P 21700, about 216 Wh | does not fit | does not fit |
| 4S3P 18650 (Samsung 35E), 144.7 Wh minimum | fits shrink-wrapped, three cells across, board P flat at its south end: 1.35 mm spare across the pocket, which is less than the case wall's own uncertainty (corrected 26 September 2026: the 1.35 mm was taken against the X 178 of appendix 32.62, which is not a Peli surface; at the worst of Peli's figures the block keeps 1.85 mm to the floor fillet and 7.38 mm to the east wall, `CASE-MARGINS.md` M4a, M4b, on the design basis only) | does not fit |
| 4S2P 21700, about 144 Wh | fits shrink-wrapped and staggered, marginal in height | does not fit |
| any of them in `pack_4s.py`'s walled box | does not fit (a three-across 18650 block needs 60.65 mm against 58) | does not fit |

So, INFERRED from the committed board heights, the pocket is expected to hold about 145 Wh at most and only without a rigid enclosure, and no pack is expected to fit the west pocket, so a second pack there is not expected to be possible with this board set.

**The owner ruled the pack on 26 September 2026 (D-06), to that finding:** one 4S3P pack of Samsung INR18650-35E cells, about 145 Wh, shrink-wrapped in the east pocket, subject to the case measurement, which the owner withdrew on 26 September 2026. Missions longer than the pack rely on vehicle or solar input. The runtime requirement is battery-only hours in the idle and typical modes at +20 C for an aged pack; the number is not computed yet, so no runtime is stated here. The owner reversed D-08 on 26 September 2026 ("you have the CAD files and all the measurements why do you need from me to measure an old case?"): no case measurement and no mock-up are asked of him. Every case-dependent margin is computed against the worst of Peli's own figures (`CASE-MARGINS.md`), and a margin that rests on a tolerance no source states is OPEN; the design targets the current moulding (D-08a), and the OPEN margins, the seals and the stack-up are shown on hardware, on a targeted unpowered mock-up in a new case of that moulding (**Corrected 27 September 2026 (MESHSAT-1357, the case set C1 to C6):** the checks of the rows that can move a board are required before the layout entry of boards A, B, E and P, which is BLOCKED on the owner's purchase decision D-09, FEA-007, `CASE-MARGINS.md` section 7 and `CASE-FIT-UNCERTAINTIES.md` sections 2 and 7; boards C, D and E5 are not held by it and the other checks run at the build; it read "for the build stage"). Two session items follow from the ruling: `pack_4s.py` is redesigned (its rigid box fits nothing), and the 4 A charge setting is lowered for cell life.

## 4. Leads

| Lead | From | To | Wire | Connector |
|---|---|---|---|---|
| Pack power (fused at the pack: the 25 A blade `F1` and, behind it, the chemical fuse `F2` of D-15) | board P's two 12 AWG leads (`W_P`, `W_N`, `gen_sch_p.py:347-348`), along the front wall | E6 `J_BATT` (XT60) | 12 AWG silicone, 350 mm | XT60 pair |
| Pack SMBus | P1 `J_SMB`: JST-XH B4B-XH-A, 1x4, 2.50 mm (1 SMBC, 2 SMBD, 3 PACK_N, 4 PRES; `gen_sch_p.py:514`, LCSC C144395, B4B-XH-A(LF)(SN), carried by the generator since round 8, R8P-02; C594232 from `lcsc_fill.py:158` was the gold -G variant JST's catalogue does not list) | E6 `J_SMB`: the same JST-XH B4B-XH-A, 1x4, 2.50 mm, in P1's pin order (1 SMBC, 2 SMBD, 3 GND, 4 PRES to the sensor controller's GPIO17; `gen_sch_e.py:218` at `45bde541`) | 26 AWG twisted, 350 mm, XH housing to XH housing, straight (pin n to pin n) | **Corrected 26 September 2026 (twice).** This row first said "XH2.5 x 6", then recorded that no lead mated both ends: E6 carried a 2.54 mm 1x6 pin header left from the withdrawn BB-2590/U, and a straight lead would have crossed clock and data. As generated since `faf8c981` both ends are the same JST-XH 1x4 in P1's order; P1's pin 3 is `PACK_N`, the pack's own negative lead, so the lead's return does not bypass the shunt; E6's sensor controller is the gauge's only SMBus host (the charger on A22 has no conductor to P1). `check_contracts.py` checks the lead as a cross-board contract since `93138ac1` (the same family, pitch and pin count, pin n's role at both ends, P1's return on its own negative lead, every SMBus clamp returning to it). |
| Vehicle and shore DC | D38999 receptacle on the back-wall plate, DC pair | E6 `J_DCIN` (JST-VH), the lead tied along the back wall, the west end wall and the front wall | 18 AWG, 500 mm | VH crimp |
| Solar | D38999 receptacle, spare pair | E6 `J_SOLAR` (JST-VH), with the DC lead | 18 AWG, 500 mm | VH crimp |
| Block signal wires | E6 `J_BLK` (twelve lands) | dock block wire lands, underside | 24 AWG, 60 mm each, named on the block's legend | soldered both ends |
| Block power pair | E6 `P_CP` and `P_CN` | dock block wire holes | 12 AWG silicone, 60 mm | soldered both ends |
| MAIN button | C7 `J_MAINSW` (two solder lands on the underside, beaded) | A22 `J_MAINSW` (XH2.5) | 24 AWG twisted | XH2.5 at the A22 end; unplugs there |
| PI button | SW_PI's contacts | C7 `J_PIJ2` lands (the panel controller reads it on U1 P1.3; nothing leaves the backer; DRAFTED by record l8r2 at `29ffb518`, PROVISIONAL until l8r2's apply_gen_sch_c_pibtn.py is released and board C regenerated; as generated no controller pin reads it, the panel firmware's F-01) | 24 AWG | soldered, beaded |
| Panel ribbon | B16 `J_PANEL` | C7 `J_PANEL` (SMD box header on the underside) | 26-way 1.27 ribbon, 350 mm | IDC 2x13 both ends |
| A to B ribbon | A22 `J_AB1` (top) | B16 `J_AB1` (underside, the same case XY) | 26-way 1.27 ribbon, 80 mm, folded once | IDC 2x13 both ends |
| Mezzanine harness (USB pair, PTT mirror, inhibit, PA rail state, I2C, 3.3 V) | A22 `J_MEZZ1` | D8 `J_HARN1` | 16-way ribbon, 60 mm | IDC 2x8 |
| Mezzanine 5 V (2 A eFuse on A22) | A22 `J_MEZZ_PWR1` (VH) | D8 `J_PWR1` (VH) | 18 AWG, 60 mm | VH |
| Slot rails, 3 x (5.1 V: AP64500 5 A bucks on slots 1 and 3, an LM5176 stage on slot 2, each INA226 monitored; `gen_sch_a.py:840-841` and `:873` at `45bde541`, corrected 26 September 2026 from "6 A converters") | A22 `J_5V_S1..3` (VH) | B16 `J_5V_S1..3` (VH) | 16 AWG, 150 mm | VH crimp both ends |
| Device rail (5.1 V, an LM5176 stage with a 7.2 A minimum limit, `gen_sch_a.py:881` at `45bde541`) | A22 `J_5V_DEV` (VH) | B16 `J_5V_DEV` (VH) | 16 AWG, 150 mm | VH crimp both ends |
| PoE feed (54 V) | A22 `J_54V` (VH) | B16 `J_54V` (VH) | 18 AWG, 150 mm | VH crimp both ends |
| PA rail (13.8 V, EMCON gated) | A22 `J_PA` (VH) | the RA30H1317M1 VCC pins on the plate | 16 AWG, 300 mm | VH at A22, soldered at the module |
| PA gate bias | D8 `J_VGG` (PH 1x2) | the module's VGG pin | 24 AWG twisted, 250 mm | PH at D8, soldered at the module |
| PA drive | D8 `J_PAIN` (U.FL) | the module's RF input pin | RG-178, 250 mm | U.FL at D8, soldered at the module |
| PA output | the module's RF output pin | D8 `J_PAOUT` (SMA) | RG-316, 250 mm, bend radius 12.5 mm | soldered at the module, SMA at D8 |
| VHF antenna | D8 `J_ANT` (SMA) | A22 `J_RF1` (VHF jack) | RG-316, 120 mm | SMA both ends |
| Headsets, 2 x | D8 `J_HS1`/`J_HS2` (PH 1x5: SPK GND MIC GND PTT) | the U-174/U jacks on the plate | 5 x 24 AWG, 300 mm | PH at D8, soldered at the jack |
| HF rail (12.0 V, EMCON gated) | A22 `J_HF` (VH) | the QMX's DC lead (2.1 mm barrel) in the lid harness | 18 AWG, 500 mm, a lead whose least bend radius is 20 or under (it is installed at R 20, the r2 tray's loop) | VH at A22; at the unit a straight 2.1 x 5.5 plug within d 18.8 and 55.4 long (r2 record) |
| QMX USB | B16 `J_QMX` (PH 1x4) | the QMX's USB-C in the lid harness | USB 2.0 lead, 500 mm, a lead whose least bend radius is 20 or under (installed at R 20) | PH at B16, USB-C at the unit, its overmold within 8.6 high, 12.35 wide and 35.4 long (r2 record) |
| HF antenna | the QMX's BNC in the lid harness | A22 `J_RF2` (HF jack) | RG-316, 500 mm, installed at R 12.5, the tree's figure for its least bend radius | BNC male at the unit within d 20.0 and 42.9 long (r2 record), SMA male at A22 |
| Monitor supply (the pack node, 14.4 V nominal, behind a 1.2 A eFuse that trips above about 17.6 to 19.0 V; corrected 26 September 2026 from "12 V") | A22 `J_MON` (VH) | the Xenarc's DC lead below the plate | the monitor's own lead, spliced under shrink | VH at A22 |
| Monitor HDMI | B16 `J_HDMI` | the Xenarc's HDMI lead | the monitor's own cable, 500 mm | HDMI A at B16 |
| Monitor touch USB (full speed, on board D's spare hub port: the session's choice SC-HF-06 of 27 September 2026, `HW-FW-CONTRACT.md` section 8, `pcb_interfaces.yaml` IF-MON; corrected from "a B16 slot hub header", which named no designator) | D8 `J_USB3` (PH 1x4: 5 V, D-, D+, GND) | the Xenarc's USB lead (a type A plug) | an adapter made up at build: a USB A receptacle to PH 1x4, 24 AWG, to the monitor's lead | PH at D8 |
| Camera | B16 `J_CAM` (PH 1x4) | the camera module behind the plate window | USB 2.0 lead, 300 mm | PH both ends |
| Ethernet | B16 `J_ETH` (RJ45) | the sealed RJ45 on the connector plate (PoE out on 1-2 and 3-6) | Cat 5e patch, 400 mm | RJ45 both ends |
| USB-C outlet, power only (D-12) | A22 `J_USBC_OUT` (5-pin: VBUS CC1 CC2 GND GND; the ESD array `U31` on CC1 and CC2, D-17, `gen_sch_a.py:1015-1026` at `45bde541`, to be placed at the header in board A's next phase) | the sealed USB-C receptacle on the connector plate | 18 AWG VBUS and GND, 26 AWG CC | soldered at the receptacle |
| USB-C outlet, data side | none since `458b2873`: the outlet carries power and CC only (owner ruling D-12) | | | **Corrected 26 September 2026 (S-07):** this row was the pigtail's data side on A22's `J_USBW`, which is now the Glenair's lead (the row below) |
| Wall USB host (console and key fill, D-12) | A22 `J_USBW` (PH 1x4: VBUS D- D+ GND; the pair `USB_WALL` from B16's bank 3 hub, port 3, over the A-B wall-port ribbon `J_AB2`; VBUS from the eFuse `U32`, 0.9142 A nominal limit (TPS2596 equation 7, SLVSET8A p.28), switched by A22's expander; `gen_sch_a.py:1668-1669` at `e57a7365`) | the Glenair 233-370 feed-through on the connector plate | USB 2.0 lead, 400 mm | PH at A22, USB-A at the feed-through. **Corrected 26 September 2026 (S-07):** this row named a B16 `J_USBX` that no generator defines, and the D-12 move it called owed is generated since `458b2873` |
| Cooler fans, 3 x | the CM5 Coolers | B16 `J_FAN1..3` (SH 1.0) | the coolers' own leads | SH housing |
| Mixer fans, 2 x | the two IP68 fans on their brackets at the stack's ends | E6 `J_FAN1`/`J_FAN2` | the fans' own leads | SH housing |
| Heater mat (a regulated 12.0 V from the buck `U33` behind the eFuse `U22`, the mat's own 12 V and 7.5 W rating, `gen_sch_a.py:1047-1076` at `45bde541`) | A22 `J_HEAT` (XH2.5) | the RS PRO 245-556 mat under the pack | the mat's PTFE leads | XH2.5 at A22 |
| Outside sensor pod | the pod on the connector plate | E6 `J_POD` (PH 1x4: 3.3 V GND SDA SCL) | the M8 receptacle's inside pigtail, 400 mm | PH at E6 |
| Sensor modules | the DCF77, Geiger and lightning boards on their standoffs beside E6 | E6 `J_DCF`, `J_GEIGER`, `J_LTG` | 3, 3 and 5 x 24 AWG, 100 mm | PH |
| Lid and tamper reed | the Littelfuse 59140 reed under the frame (its 57140 magnet in the lid) | E6 `J_TAMP` (JST-XH 1x2, `gen_sch_e.py:524-542` at `45bde541`) | the reed's own 1000 mm leads | XH at E6; added 26 September 2026 (S-07) |
| Water electrodes | E6 `PAD_W1`/`PAD_W2` | two bare copper strips on the floor at the low corner | 22 AWG, 150 mm | soldered |
| GNSS, LoRa pigtails | B16 `J_GNSS1`, `J_LORA1` (U.FL) | A22 `J_RF4`, `J_RF11` | U.FL to SMA, RG-178, 150 mm | U.FL at B16, SMA at A22 |
| WiFi link card pigtails, 4 x | the two AW7915-AED cards' MHF4 connectors | B16's changeover inputs `J_W1A`, `J_W1B` (slot 1 card) and `J_W3A`, `J_W3B` (slot 3 card) | MHF4 to U.FL | both ends pushed on |
| WiFi link antenna pigtails, 2 x | B16's changeover outputs `J_WOA`, `J_WOB` (U.FL; two SKY13351 switches move both antennas to the slot 3 card under the voted changeover, `gen_sch_b.py:1253-1272` at `45bde541`) | A22 `J_RF6`, `J_RF7` (P2P A, P2P B) | U.FL to SMA, 200 mm | U.FL at B16, SMA at A22; corrected 26 September 2026 (S-07) from one card wired straight to A22 |
| 5G pigtails, 2 x (a third, ANT3, when D-07's third jack reaches A22) | the RM520N-GL's ANT0 and ANT2 receptacles (the module has no MAIN or DIV port) | A22 `J_RF8`, `J_RF9` (legends 5G MAIN and 5G DIV) | MHF4 to SMA, 200 mm | MHF4 at the module, SMA at A22 |
| Iridium | the RockBLOCK 9704's SMA | A22 `J_RF10` | RG-316, 120 mm | SMA both ends |
| SDR | the LimeSDR Mini's SMA | A22 `J_RF5` | RG-316, 150 mm | SMA both ends |
| WiFi 2.4 | one Compute Module's antenna-kit lead (slot 1) | A22 `J_RF3` | the kit's own lead (U.FL to SMA) | SMA at A22 |
| RF jumpers, 11 x | the float clamps on E6 (Radiall R222M80500 right-angle plugs, crimped, tied into the clamp) | **Corrected 27 September 2026 (MESHSAT-1357, the case set C1 to C6):** the inner jacks of the PolyPhaser GTH-SFF-AL arrestors on the RF entry plates (C2, C4): west VHF, HF, WIFI 2.4, GNSS, SDR, WIFI P2P A, WIFI P2P B at Y -93, -62, -31, 0, +31, +62, +93; east 5G MAIN, 5G DIV, 5G ANT3, IRIDIUM, LORA at Y -62, -31, 0, +31, +62; all at Z 59. Until 27 September 2026: eleven Amphenol 132170 couplers at Z 88 | RG-316, each cut to its route plus 20 mm, 252 to 432 mm (`CASE-MARGINS.md` 3.4; it read 150 to 250), bend radius 12.5 mm | SMP-MAX plug at the clamp, right-angle SMA male crimp plug at the jack (the pick is OPEN: M17g and M17x) |
| Connector plate | **Corrected 27 September 2026 (MESHSAT-1357, the case set C1 to C6):** 114.0 x 68.3 x 5.0 aluminium (C3, `v2/release/case-2026-09-27/connector-plate/`); until 27 September 2026 54 x 82 x 3 between ribs | the back long wall (hinge side) between the hinge fairings, centred at X 0, Z 18.3 to 86.6 | six M4 x 25 A2 at X +-51.1, Z 24.2, 50.1 and 76.0, a bonded sealing washer under each outside head, a plain washer and a Nyloc inside, in a cross pattern; 2 mm closed-cell gasket | carries all six ruled items at the centres of `CASE-MARGINS.md` 3.3: A the sealed RJ45 (-28.5, 36.6; pick OPEN, the PX0833 fails the shell 15 envelope and 54 V), C the D38999/20 shell 13 DC receptacle (+4.2, 34.0), B the sealed USB-C (+33.7, 36.6; the PXP4043/C panel drawing OPEN), E the pod over its M8 receptacle (-30.0, 70.0; sheet not held), D the 233-370 USB feed-through (+4.6, 67.0), F the M6 ground stud (+34.6, 64.5); A, C and D each on a Glenair 930-001 gasket with M3 into threads tapped in the plate. The OPEN picks' cut-outs are PROVISIONAL (red on sheet 3) |

Every lead tied at both ends; the rod stack's edge carries the vertical runs with a tie base per bay; the lid harness (QMX USB, 12 V, BNC jumper) has a service loop at the hinge.

**External cables (appendix 32.32, sheets in `vendor/d38999/`).** Two cables leave the case through the connector plate on the back wall.

| Cable | Kit end | Cable | Far end |
|---|---|---|---|
| DC lead | Glenair D38999/26FC4SN plug (shell 13, insert 13-4, four M39029/56-352 size 16 socket contacts, key N, electroless nickel), crimped with the M22520/1-01 tool and the M22520/1-04 positioner, seated with M81969/14-03; Glenair M85049/38S13N self-locking straight strain relief on the plug's M18 x 1 thread | Lapp OLFLEX ROBUST 210 4 x 1.0 (article 0021917, 6.6 mm, TPE, outdoor), or Alpha Wire 25064 (18 AWG 4C, TPU, 6.58 mm); 2 m | the four cores split under adhesive-lined shrink into two 0.3 m tails: the DC pair to the shore supply or to the NATO 2-pin vehicle plug (9 to 36 V, the front end takes either), the solar pair to the panel |
| USB host lead | Glenair 233-340 plug (shell 15, USB 2.0 Type A male front and Type A female back, key N, horizontal, with the 770-028 shrink boot), screwed onto the feed-through | a standard USB 2.0 Type A male to Type A female extension, 1.5 m, its plug in the back of the 233-340 and the boot shrunk over its jacket | the extension's Type A female, into which the device's own lead plugs |

Contact assignment of the DC plug: A DC positive, B DC return, C solar positive, D solar return; Lapp cores 1 to 4 in that order, Alpha colours black, red, white, green. The cable's insulated cores must lie inside the size 16 grommet window of 1.65 to 2.77 mm (MIL-DTL-38999 Table IV); the Alpha cores are 2.0 mm, the Lapp core diameter is measured on the reel before that cable is used.

The dock interface is not a lead but belongs in the same reading. Twelve Preci-Dip 813 contacts in `J_DOCK` on A22's underside land on the raised block's targets: pins 1 to 7 ground, 8 `SHORE_INHIBIT`, 9 and 10 the USB pair of E6's sensor controller, 11 ground and 12 the hot stop line HOT-R1 (`DOCK_SPARE`, since stream w4ae), with `VIN_RAW` (the 9 to 36 V input and the solar tracker's output, passed up to A22's front end) on four 9 A spring pins of its own, `J_VR1` to `J_VR4`, with its return on four more, `J_VN1` to `J_VN4`, since EQ-16 (`gen_sch_a.py:294` and `gen_sch_e.py:660` at `e57a7365`; at `45bde541`, `gen_sch_a.py:225` and `gen_sch_e.py:488`, pins 1 to 4 carried `VIN_RAW`; corrected 26 September 2026, S-07: this sentence put the wall outlet's console pair on 9 and 10). Beside them, nine Mill-Max 0858 class pins carry the pack current: four on the node, four on the return, and one longer pre-charge pin that mates first through a 10 ohm resistor so the converters' input capacitance does not draw an arc across the main pins. The eleven RF joints mate at the same time, and the whole set parts when the stack is lifted.

## 5. Conformal coating

IPC-CC-830 acrylic (MG Chemicals 422B or equal) on A22, B16, D8, the dock strip E6 and the dock block E5 after the bench fit, two thin coats. Masks (kapton) before coating: every connector face and its keying, the spring-pin targets and the pack targets on E5 and the pins on A22, the SMP-MAX receptacles and the SMA and U.FL bodies, the six Compute Module receptacles and the seven M.2 sockets (assembled cards are not coated), the RockBLOCK bracket, the LimeSDR receptacle, the SA868 module and the relay, the water electrodes and the sensor headers on E6, the test points that the bench list uses. C7: the whole underside is coated after the silicone beads have cured, with `J_PANEL`, `J_EPD`, the lead lands and the eight standoff rings masked (the rings bond the backer to the plate); the top side is not coated where the LEDs stand. The plate is bare anodised aluminium.

## 6. Labels (MIL-STD-130 style)

- Plate nameplate field at `NAMEPLATE` (78, -101), 76 x 26: "MESHSAT FIELD KIT", P/N MSK-FK-1450, S/N, REV A, a 10 x 10 mm data matrix with the S/N, "MADE IN NL"; laser-marked with the plate's other legends (`v2/cad/face_plate.py`).
- Every board: P/N, S/N, REV silk fields near the title block silk.
- Case: asset label in Peli's label recess; "RF HAZARD DURING TX" 20 x 40 mm next to the VHF arrestor; the bulkhead legend strips beside the arrestor rows (**Corrected 27 September 2026 (MESHSAT-1357, the case set C1 to C6):** west VHF HF WIFI 2.4 GNSS SDR P2P A P2P B, east 5G MAIN 5G DIV 5G ANT3 IRIDIUM LORA, C2).

## 7. Removal and refit

Open the lid (the QMX tray swings with it; unplug the lid harness at B16 `J_QMX`, A22 `J_HF` and `J_RF2` if the lid is to come off its hinge; the QMX itself comes out of the r2 tray by its three plugs, the frame's six screws and the frame), take out the ten plate screws, lift the face plate with the backer C7, the monitor, the PA module and the switches hanging under it (the panel ribbon, the MAIN lead, the headset pigtails, the PA leads and the monitor's three leads unplug at the B16, A22 and D8 ends), then lift the A22 + D8 + B16 stack straight up through the frame window (349.65 x 233.83; A22 is 240 x 160, B16 330 x 200; 8.25 mm per side at the worst, `CASE-MARGINS.md` M7). **Corrected 27 September 2026 (MESHSAT-1357, the case set C1 to C6):** the frame and its four setting legs stay in the case; the ten plate screws are 6-32 from above. No connector is unscrewed: the eleven RF joints, the twelve signal contacts and the nine power pins all part as the stack rises. The pack lifts out of its cradle after its XT60 and SMBus are unplugged at E6. Refit in reverse; the rods through the dock strip's holes align everything, and the pre-charge pin meets its target before the four main ones.

**The stack is never lifted live (owner ruling of 26 September 2026, D-14).** The dock carries `VIN_RAW` (up to 36 V) on four spring contacts and the pack node (up to 16.8 V and about 18 A) on four power pins (W3-F09), and it parts and mates whenever the stack is lifted, which leaves the E5 targets exposed at the floor. Before the stack is lifted, in this order: (1) the kit off at MAIN; (2) the vehicle, shore and solar leads unplugged at the connector plate outside; (3) the pack's XT60 unplugged at E6 `J_BATT`. `J_BATT` sits at the strip's front west corner in the case frame (`gen_pcb_e3.py:60` and `v2/cad/render/scene.py:269`, X -138, Y -108); whether a hand reaches it with the stack in place has not been checked against A22's and B16's outlines or in the owner's case, and if it does not, an in-line disconnect on the pack lead is a session item. While the stack is out, an insulating cap goes over the E5 block, and it comes off only when the stack is about to go back. Lifting with the pack connected is an accepted and recorded residual risk; a hardware "stack present" interlock on the spare dock contact is studied at Review D, because it touches the pack protection of decision 40. The insulating cap is not yet drawn or sourced.

## 8. Commissioning after assembly

`TEST-PLAN.md` is the qualification programme; the list below is what to check once, in this order, on the first kit.

1. Dock strip alone: the 20 V bus at the block lands with 9, 12, 24 and 36 V in; reverse polarity applied for 10 s (no damage, no output); the fuse blows on a bolted short. Then the tracker: a panel or a bench supply through a series resistor, and the tracking point holds while the load changes. The sensor controller enumerates on the bench USB lead and reports every sensor it has.
2. Dock block alone, before the stack goes on: continuity from every wire land to its target, and no continuity between neighbours. This is the last moment the lands are reachable.
3. A22 alone, pack not connected: a bench supply at 14.4 V on the node contacts through a 5 A limit. Each rail comes up at its own converter (the three slot rails and the device rail at 5.1 V within 0.1 V, the PA rail at 13.8 V, the HF rail at 12.0 V, the PoE rail at 54 V, the 3.3 V logic); 3 A drawn from a slot rail holds it above 5.0 V. The charger enumerates on the bus, the monitors read, and the main power control turns the rails off and on from the MAIN button. With `EMCON_HW` low the PA and HF rails stay off (corrected 26 September 2026: this read "high"; the line is active low; since board A's round 8 `PA_EN` = `TX_INHIBIT_n` AND `EMCON_HW` AND `PA_HOLD` in `U35` and `U36`, and `HF_EN` likewise in `U37` and `U38` (`gen_sch_a.py:1572-1575` at `e57a7365`), and with the ribbon out `R102` pulls `EMCON_HW` low and `R145` pulls `TX_INHIBIT_n` low (`:1597-1598` at `e57a7365`), so on a bare A22 the two rails stay off until both lines are driven high).
4. Charge: 12.0 V on the DC inlet, the pack connected with its SMBus. The charger delivers into the pack the current the panel controller programmed, and the pack's gauge (BQ4050) opens its own charge FET when its cell-surface thermistor reads outside 0 to 45 C (`pcb_pack_protection.yaml` CHARGE_TEMPERATURE_WINDOW). **Corrected 26 September 2026:** the step read as if the charger saw the thermistor, and the BQ25731 has no thermistor input (TI SLUSE66A, Table 7-1). Since `faf8c981` and `458b2873` the charger's cell-count strap selects 4S and the SMBus lead mates (`PANEL.md` section 10, section 4 above); the kit's loads sit on the charger's system side, so read the pack's own current at the gauge rather than the charger's input current (corrected 26 September 2026, S-07: this step said it could not pass).
5. The stack with B16: each module boots from its rail with the other two slots disabled, then all three together; every USB device enumerates on its hub; the Ethernet switch links all three and the wall port. Record each rail's current at idle and with the display on.
6. Bursts: 5G registration, one Iridium session, one LoRa transmission and one VHF key-down in turn, each rail watched at its connector, then all within the same second: what is being recorded is the margin.
7. Panel: the panel controller enumerates; lamp test lights all seventeen controller-lit indicators (the sixteen panel LEDs `D1` to `D16`, the TX lamp `D3` among them through its tie `D17`, and the PI button's ring; `PANEL.md` section 9); BLACKOUT kills the rail; the EMCON toggle locked closed keeps the SA868 and the PA in receive while the bridge asserts PTT and opens every transmitter rail gate, and every other radio goes dark (D-05, `PANEL.md` section 6), measured with an external receiver; ZEROIZE armed shows on the e-paper and, held 5 s, performs the erase of `PANEL.md` section 6 (decision 30: the secure element's wrapping key destroyed, the running modules' RAM keys dropped, the slots cut), after which no drive unlocks; SOS closed 2 s under EMCON queues its message and tells the operator (D-10, `PANEL.md` section 9).
8. Power loss: pull the DC lead and confirm the kit keeps running from the pack and the panel shows SHORE off.
9. Shore inhibit: `SHORE_INHIBIT` high holds the front end off within a second, low restores it.
10. PA: key-downs of at most 60 s each at 30 W into a load, at least 2 s apart, each started only inside K2 and ended by C4 (`feasibility/POWER-THERMAL.md` sections 7.2 and 9.3), as `TEST-PLAN.md` T-H3 runs them; the flange sensor and a thermocouple beside it logged, and the case skin temperature recorded, the fans running. **Corrected 27 September 2026 (Review A of layer 2, finding B6; `CONOPS.md` section 4d):** this step was ten minutes of key-down at 30 W, which K1 forbids: one 60 s key-down at 45 W of heat from a +50 C plate already puts the flange at about 95 C on the record's own figure, against the RA30H1317M1's +100 C case maximum and its 90 C advice (PWR-F15).
11. Blind-mate: lift the stack and set it back three times, each time by the procedure of section 7 (kit off, outside leads and pack unplugged, the cap on E5 while it is out). Every RF path still passes, the pre-charge pin still mates first, and nothing on the block is scored.
12. Pack gauge data flash (decision 40, owner ruling of 26 September 2026), before the pack is first charged or discharged: read the BQ4050's protection thresholds and enabled protections back and compare them with `pcb_pack_protection.yaml`. Board P's second level covers cell under-voltage in hardware since `faf8c981` (D-15's first branch), so the read-back is the check D-15 keeps; only after it passes is the chemical fuse armed by closing `JP1` (`gen_sch_p.py` docstring and `:476`; corrected 26 September 2026, S-07).

## 9. Bench-fit lists (hand-fitted parts per board, not on the JLC BOM)

- A22: the Preci-Dip 813-S1-012-10-016101 spring connector and the seventeen Mill-Max 0858 class power pins on the underside (nine for the pack and, since EQ-16, eight for the input, section 4) (tails soldered on the top face), the eleven Radiall R222M00720 blind-mate receptacles, the Keystone 3568 holder with its 25 A mini blade, the inductors that have no assembler equivalent (read the ORDER-NOTES), the rail leads, the PA, HF, monitor and heater leads, the MAIN button lead, the wall USB-C leads.
- B16: the three Compute Modules (CM5108064) on their receptacles and standoffs, the three coolers with their fan leads, the two WiFi link cards (`J_M2C1`, `J_M2C3`), the 5G module with its two SIMs, the three NVMe drives, the LimeSDR, the RockBLOCK on its bracket, the CR2032, the rail and PoE leads from A22, the antenna pigtails, the HDMI cable, the camera and QMX leads, the panel and A-B ribbons; the LG290P, the E22 and the two E72 are assembled where JLCPCB stocks them, else hand-soldered.
- C7 (the backer under the plate; the switches, the jacks, the camera and the sounder mount in the plate and only their leads reach the board): the seventeen 3 mm LEDs (`D1` to `D16` and, since board C's round 8, the hardware EMCON lamp `D22`) standing on the top face under the light guides (beaded to 5.3 mm), the Floyd Bell sounder with its gasket, the three C&K switches, the NKK toggle, the three APEM toggles with their covers, the two U-174/U jacks, the camera module, the PDi e-paper on its ZIF, the RP2040 and its flash if JLCPCB has no stock, the two XH leads.
- D8: the SA868 module where JLCPCB has no stock, the G6K relay if short, the U.FL and SMA leads to the PA and the antenna, the two headset pigtails, the VGG lead; the PA module itself is a plate part.
- E6: the three Keystone holders with their blades, the JST-VH DC and solar leads, the XT60 counterpart and the SMBus socket (JST-XH 1x4), the lid and tamper reed on `J_TAMP`, the twelve signal wires and the 12 AWG pair up to the block, the printed float clamp bar (`v2/cad/float_clamp.py`: one part, twelve 8.5 mm cavities, 22 M3 x 8 into the strip's clamp holes at the mid-pitch points between cavities, each plug's cable laid in its own slot to the south or north and tied through the bar's two tie slots beside it) with their Radiall R222M80500 plugs, the DCF77, Geiger and lightning modules on standoffs beside the strip, the two mixer fans, the water strips, four VHB pads.
- P1 (inside the pack): the 25 A blade in F1, the four 2.5 mm2 solder lands (the block's B+ and B- straps, the pack's two 12 AWG leads), the five tap wires into J_CELL, the four cell thermistors into J_TS and the second level's own thermistor into J_TS2 (on the hottest cell), the SMBus lead into J_SMB; the gauge's golden image from bqStudio over the SMBus before the lid goes on, and the arming jumper JP1 left open until section 8 step 12 (corrected 26 September 2026, S-07).
- E5: nothing is placed on it by the assembler. It goes on four M3 x 6 standoffs above the strip, and the twelve signal wires and the 12 AWG pair are soldered into its plated lands from below before the stack is fitted.
- Case and face (**Corrected 27 September 2026 (MESHSAT-1357, the case set C1 to C6):** C1 to C6): the four setting legs with their VHB 5952 pads, the printed locator and the two pairs of printed wedges; the connector plate (114.0 x 68.3 x 5.0) and its gasket with its receptacles on the back wall, each on a Glenair 930-001 silicone flange gasket, the six M4 x 25 plate screws with bonded sealing washers; the twelve PolyPhaser GTH-SFF-AL arrestors on the two 6.0 mm RF entry plates with their two gaskets and sixteen M4 x 12 ISO 7380 screws on rubber-faced sealing washers (in place of the eleven Amphenol 132170 couplers at Z 88); the sensor pod on its M8; ten 6-32 UNC x 1/2 in A2 pan heads for the plate (in place of the M3 x 10 with star washers); the face seals and hardware of `vendor/seals/` and `vendor/mentor/`: the e-paper tape frames from `face-plate.dxf` (the PORON ring is dropped, C1), the 2.0 mm UV polycarbonate lens with 3M Primer 94, three Silex GP60 silicone washers, the NKK AT516 spare O-ring and AT428H boot, the APEM K seals, the Floyd Bell 61663 gasket, sixteen Mentor 1282.5004 light guides, eight PEM SO-M3-10 standoffs and two S-M3 nuts, the Xenarc window gasket, DOWSIL 3145 clear for the beads, MG Chemicals 422B for the backer's underside, the 3M 7871EC serial label; the QMX tray r2 (the printed tray and retaining frame, the 5052 lid plate, ten M3 x 5 countersunk A2, six M3 x 10 button head A2 with six M3 square nuts, two PORON 4701-30 pads, DP8005 for the plate, bonded tie mounts for the lid harness).

## Disassembly and reassembly in pictures (render set eight, 7 Sep 2026)

**Corrected 27 September 2026 (MESHSAT-1357, the case set C1 to C6):** the render set shows the superseded arrangement (the face plate under the frame's ring on M3, eleven couplers at Z 88, the old connector plate) and is not regenerated (`v2/cad/README.md`: the render scene is superseded for measurement); the sequence below stands, with the frame and its legs staying in the case and the plate's ten screws being 6-32 from above.

The concept set `v2/images/concept-1450/` carries the sequence a technician follows; every removed part is set down beside the case in the picture:

1. `meshsat-1450-assembly-1-closed.png`: the kit closed, latches shut, antennas off, cables out.
2. `meshsat-1450-assembly-2-lid-open.png`: lid open; the face plate with the monitor, the switches, the headset jacks and the e-paper is the first thing seen, the QMX tray on the lid's inner face.
3. `meshsat-1450-assembly-3-plate-off.png`: the ten M3 screws out, the face plate assembly (plate, backer C7, monitor, PA module, switches, jacks, e-paper) lifted on its ribbon and set down east of the case.
4. `meshsat-1450-assembly-4-stack-out.png`: the A22 + D8 + B16 rod stack lifted straight up off the dock's blind-mate joint (no cable unscrewed: every antenna path mates at the dock strip) and set down west of the case.
5. `meshsat-1450-assembly-5-dock.png`: the empty case: the dock strip E6 with its eleven float clamps and the pigtails from the end-wall couplers, the block E5, the sensor modules, the connector plate leads.

The pack appears as a stand-in box in the east pocket (its enclosure is not drawn yet, appendix 32.62). Reassembly is the same sequence in reverse: the rod stack lowered onto the dock (the float clamps align the SMP-MAX plugs), the face plate onto the frame and its ten screws, lid closed. Nothing has been built; the pictures are the design intent.

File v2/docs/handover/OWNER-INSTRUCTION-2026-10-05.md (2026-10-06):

# The owner's instructions of 5 October 2026: the recovery review, the 160 C correction, the review of the 13:55 report, and the P0 instruction with its two plan reviews

Filed as received (MESHSAT-1357), byte for byte inside each part below, including the owner's own typography (the saved copies'
one-line filing headers removed; the texts themselves untouched). Nothing here is edited. Parts 1 to 11 are in
`OWNER-INSTRUCTION-2026-10-04.md`. The live plan that applies these parts is `v2/docs/EXECUTION-PLAN.md`, entry of 5 October 2026
14:48 CEST; the compact blocker list part 15 asks for is `v2/docs/records/l4close/P0-POWER-LIST.md`. Part 15 made Layer 4's power architecture the only active layer; part 19 narrows that: the
deliverable is the desk engineering package for a receiving company, each layer accepted at its DESK gate in order, with physical
qualification and fabrication release as separate gates and the supplier's validation scope written down, not awaited. Prototype framing: nothing is built, bought or measured.

| Part | Received | sha256 of the part's text |
|---|---|---|
| 12. Review of the morning's recovery: the CAN fault phrase clarified (an open defect if over the limit, else the applicable requirement named) | 5 October 2026, about 10:30 CEST | `f6afeceae0c19ea7d50d9ad686288cfd1958eb3208f02e3640588518680880d7` |
| 13. Correction: 160 C typical shutdown is not a permitted temperature limit (125 C the criterion, 150 C the absolute maximum, 176.3 C a model result that fails) | 5 October 2026, about 11:00 CEST | `1d2391b5b8bf3de31d85c4193ce833f02c7abec488e1e6056eec6314ee83e493` |
| 14. Review of the 13:55 status report: continue under three workers; T11 states apart; firmware escalation not assumed; copper comparison with quoted or estimated cost; F13, F16, F17 not corrected; set 30's bounded scope | 5 October 2026, about 14:05 CEST | `d7aadb430e574c733b3afff675005b76298d3d94ee0bf07c834e16dd3cb00268` |
| 15. P0 power closure and strict layer-by-layer execution (supersedes the permission to keep later layers moving; stop and preserve; one connected power correction with three workers; the Layer 4 exit gate; convergence; layer order; checkpoints) | 5 October 2026, 14:20 CEST | `91c55cc21c8152c33213b2938330d8ebd874a08b035b0f55de7f381a909c5bee` |
| 16. Review of the P0 execution plan: proceed after four targeted amendments (calibration and layout bounds need a feasibility basis; the integration order and one combined base; preserve work and start engineering beside the clerical work; the external closure path made actionable) | 5 October 2026, about 14:45 CEST | `a80ab901ae447f789bc74ec0cfbfc0103725c44d73c4282764908d02c489f726` |
| 17. Second review of the revised plan: READY to approve for execution; the baseline watchpoint; 14 to 18 h is a desk candidate, not Layer 4's closure | 5 October 2026, about 14:55 CEST | `14f5dcc8fc2aacc4a5a9e33a06b321021651889cf5d7b6dfeee12bc3776d8b8d` |
| 18. Review of P0 checkpoint 1: continue the authors; finish the external decision packet (U-02's per-mode reconciliation and the mock-up's sum, U-04's evidence route apart from the whole-kit release, U-01's two kinds of evidence) | 5 October 2026, about 15:30 CEST | `62351f9c8ca4a11b1328b5fcfb161c680b17701335242d8a3d505b5c900085a2` |
| 19. Handover scope amendment and review of the external packet: the deliverable is the desk engineering package for a receiving company; sequential DESK acceptance per layer; the packet reframed as the supplier validation annex with three corrections (a failed arrangement is not a requirements conflict; the mock-up sum; investigating the Saft option apart from adopting it) | 5 October 2026, about 15:45 CEST | `d448616ce3607d9653fe47efea771aa9a68e31198ec943bf52a9f4bf8262b02a` |
| 20. Targeted revision check of the supplier annex: its revised scope accepted (not the circuitry); two follow-throughs (residual owner-role wording; the live plan must show sequential desk-handover gates governing while the design and fabrication gates stay honest) | 5 October 2026, about 15:58 CEST | `0755be17a7931895b431c0d75419d15246c46e1d9e9c88554b31aa58927f539d` |
| 21. Targeted review of P0 checkpoint 2: continue; the independent check of T10's drafted correction must establish four things (the air and tolerances, the CAN service under the share, enforceability, the match to C-DEV rev 2); F01's next selection record disposes of cx44's ten findings individually; the freed checker slot on P0-7 is within the limit | 5 October 2026, about 16:08 CEST | `9db73b773db19c04c5306dbdaafc885e96a522362adbb2fa7663a252c8f05131` |
| 22. Targeted review of P0 checkpoint 3: continue; the guard's latent-fault disposition (L8P-D9) needs an engineering basis per fault or the defect stays open with a correction; the 146.4 C babbling-supervisor case needs its applicable criterion named (125 C design criterion kept distinct from the 150 C absolute maximum); revision V tied to the part specification, sourcing and case selection; F01 and the solar alternative provisional until checked | 5 October 2026, about 17:05 CEST | `9dbcee0e973b2401387a7a68e7a2e869c2b1cfa70b861bfb3907c6e91580c275` |
| 23. Review of P0 checkpoint 4: continue; D-10 and S1 are unresolved protection engineering (the model reports voltage over the 80 V row), carried as a remaining-engineering item with the failing cases, the requirement per case, the correction route and the provisional outputs; B2 an unapproved partial interface proposal whose cold-connection guarantee cx45 verifies; R602's final margins on the connected candidate | 5 October 2026, about 17:50 CEST | `5ec043b65723f51bf0bd1f7923af801abc84f1ba176d3952b83e3f4531197faa` |
| 24. Review of P0 checkpoints 5 and 6: the candidate NOT CONFIRMED; finish the bounded correction round and cx46 (cx45's findings the before/after checklist; a diagnostic's bounded interval covers faults after start-up and in the diagnostic itself; the governing inputs in the candidate); the latent-guard owner question superseded; B2 optional; an unsupported correction is handed over as remaining engineering, never as qualification-only; desk-handover readiness assessed apart from power closure and fabrication release | 5 October 2026, about 19:15 CEST | `1872d381fa5a9acc22da3049331cc9a052a51cd8eb4a90ecfac29ecc14d28bfe` |
| 25. Review of P0 checkpoint 7: continue to cx46; B2 unselected and withdrawn as drafted, no longer an owner action, the approved interface retained; cx46 to judge whether the handed-over guard and CAN cases weaken any protection, thermal or service bound; the integration gate binds the reviewed and the integrated revisions with the intervening changes classified | 5 October 2026, about 20:10 CEST | `3d7a893368c91aec176f57b7e4dbc39a24e4710c378d7d26a6e5f2cb6c9417a0` |
| 26. The MeshSat communications bootstrap: a durable request/reply channel between the owner's supervisory review session (through its Codex tunnel) and the engineering coordinator, with the roles preserved, a minimal request/ACK/result protocol, a transport-only continuation pointer on the runner, a genuine round-trip test, and the engineering state untouched (public copy: host, path, session and tunnel identifiers replaced by placeholders; the sha256 is of the verbatim text kept on the runner) | 5 October 2026, about 21:40 CEST | `6840bbc8ad1d056cc8c95f523b4f30047755457d0e63aaaccc661d737cc9b136` |

---

## 12. Review of the morning's recovery: the CAN fault phrase clarified (an open defect if over the limit, else the applicable requirement named) (as received)

**The reported recovery looks properly controlled:** staged work is backed up, three authors resumed from checkpoints, and the rented boxes are stopped with disks retained. No new broad prompt is needed.

One phrase needs clarification in Slot C’s report: **“junction temperatures under CAN-bus faults, outside the criterion.”**

- If temperatures **exceed the permitted limit**, retain an open defect.
- If the fault case is **outside T10’s scope**, identify the applicable requirement and where that case is handled.

The 4.18 V pre-regulator remains a drafted candidate until checked. The next useful milestones are Slot C’s completed report and V5’s firmware verdict.

---

## 13. Correction: 160 C typical shutdown is not a permitted temperature limit (125 C the criterion, 150 C the absolute maximum, 176.3 C a model result that fails) (as received)

**One correction: 160 °C typical shutdown must not be treated as a permitted temperature limit.**

Keep these separate:

- **125 °C:** T10’s stated design criterion.
- **150 °C:** the manufacturer’s absolute maximum junction temperature—not an operating target.
- **160 °C typical:** shutdown behavior, with no guaranteed maximum trip temperature stated. It cannot prove protection below the absolute maximum. [diodes.com](https://www.diodes.com/assets/Datasheets/AP2112.pdf?utm_source=chatgpt.com)

The reported **176.3 °C is a model result**, not a measured temperature. It fails the stated thermal bounds; the real device might shut down or cycle, but that does not establish acceptable fault behavior.

Claude should retain the applicable fault finding until a supported correction or protective response meets the required temperature and service criteria. This clarification can join the current author’s work.

---

## 14. Review of the 13:55 status report: continue under three workers; T11 states apart; firmware escalation not assumed; copper comparison with quoted or estimated cost; F13, F16, F17 not corrected; set 30's bounded scope (as received)

(The owner's review of the 5 October 13:55 status report, as pasted in the session at about 14:00 CEST; full text kept in the session
log's source. Its continuation prompt, binding:)

Continue the current work under the three-worker limit; do not restart it or add another broad review.

Finish V5F, V2RG and V6 against their actual candidate revisions. Report active versus queued jobs accurately, and preserve every review verdict. Then define and execute set 30's bounded integration scope under the existing gates, with explicit open and conditional items. Give the candidate, remaining prerequisites and next completion checkpoint.

Make these small reporting/decision corrections in the normal update:
- T11: distinguish research delivered, review corrections open and three-radio fit not demonstrated. Provide the plan, Astra's recheck and O-1a–O-7 table for the SDR decision. A one-radio pilot is not approval of the final architecture.
- Firmware escalation: do not assume an engaged supplier firmware engineer. If escalation becomes necessary, preserve the reproducer and unresolved defect, specify the capability needed and identify who must secure it. A review limit does not close a software defect.
- Copper: finish the viable-options comparison with technical basis, recommendation and quoted or explicitly estimated cost; disclose any pricing unknown.
- Keep CAN fault findings F13/F16/F17 out of the list of corrected defects while they remain open.

No new purchase, vendor contact or requirement change is authorised by this clarification. Continue all independently eligible layer work and keep fabrication release blocked until its own criteria are met.

---

## 15. P0 power closure and strict layer-by-layer execution (supersedes the permission to keep later layers moving; stop and preserve; one connected power correction with three workers; the Layer 4 exit gate; convergence; layer order; checkpoints) (as received)

# Owner instruction: P0 power closure and strict layer-by-layer execution

This instruction supersedes earlier permission to keep later layers moving, fill spare worker slots with unrelated tasks, or leave current workers running because they are busy. Preserve existing work and evidence. Change the execution priority now.

Prepare a short executable plan, then execute it through the normal plan-mode handoff. Do not respond with another general constitution or research programme. My objective is the earliest defensible completion of the power architecture, followed by each remaining layer in order. P0 is the execution priority; retain the actual engineering severity of each finding separately.

## 1. Stop the current allocation and preserve the work

- Interrupt all currently assigned Claude and Codex/Astra workers. Cancel their current assignments and queued continuations, including SDR research and unrelated firmware, mechanical, component and documentation work. Do not wait for their current rounds to finish.
- Capture each branch tip, staged and unstaged changes, relevant untracked files, logs, and a short resume note. Preserve incomplete work explicitly as incomplete. If an agent cannot respond, the coordinator captures its worktree.
- Stop project-owned child jobs and monitors that would continue these assignments. Preserve partial outputs separately from previously valid outputs. Do not kill unrelated processes, discard changes, reset branches, delete worktrees or overwrite accepted evidence.
- Verify that no stopped assignment can continue writing or relaunch itself. Report any process you cannot stop and what it can affect. Target a brief recovery checkpoint, not an hour of packaging.
- Stop rented compute that is no longer useful; retain disks and prepared environments. Nothing is destroyed. Existing compute spending authority remains; hardware purchases and external messages remain subject to their existing authorisation boundaries.

If active plan-mode restrictions prevent these actions, state that they have not happened, identify what remains running, and make this the first execution step. Do not claim workers are stopped merely because a plan says to stop them.

## 2. Establish the current baseline and the actual power blockers

Read the owner brief, accepted requirements, current main, and the latest relevant branches and review records. The 13:55 report named main `aa32332c`; verify the live state rather than assuming it remains current. Preserve already supported corrections instead of repeating their derivation without cause.

Use the existing findings register. Produce one compact current list with: finding, failing operating/fault case, requirement or limit, correction needed, owner, evidence needed, dependency and closure test. Distinguish:

1. A desk-fixable circuit, calculation, firmware/protection or interface defect.
2. Missing evidence that can still be obtained or bounded at the desk.
3. A genuine external dependency: a manufacturer statement, measurement, supplier engagement or owner decision.

Start with the remaining power defects, including F01/all-transmit, CAN fault findings F13/F16/F17, I-03 and its ground return, T10, eFuse settings and their coupled protection/thermal effects. Check the current disposition of solar protection, battery FET sharing, thermal protection and coupon-method findings. Do not reopen corrected items merely because their identifiers occur in old reviews; do not omit an open item because it belongs to another layer's record.

F01 must receive an author and a next engineering action immediately. It must not remain undrafted while all available slots work on secondary reporting or review tasks.

## 3. Keep the approved requirements fixed

Retain the current owner-approved baseline: internal battery and solar, no external battery, HF and tablet retained, the approved enclosure and pack ruling, optional tablet charging, and the 48–72-hour runtime objective correctly distinguished from mandatory service.

Use the exact repository requirements for all-transmit operation, starting voltage, fans, compute loads, source windows, temperature modes and fault service. Retain REQ-016's approved solar window. Do not solve a mandatory power defect by silently raising the operating floor, reducing service, turning off required fans, relying on typical compute consumption in a different case, or changing thermal requirements.

The three-SDR proposal is paused and unadopted. Keep its loads and fit assumptions separate from the approved baseline. Preserve the study for a later owner decision.

Leave Layers 1–3 accepted unless a specific, evidenced contradiction actually requires an amendment. If a change of requirement, pack, enclosure, service or spending authority becomes necessary, present the smallest concrete decision with consequences. Do not make that change yourself or conceal it in an engineering assumption.

## 4. One connected power correction, with three workers maximum

The coordinator remains accountable for convergence and integration. Assign fresh, bounded briefs using the recovered work:

| Slot | Responsibility |
|---|---|
| A | One power-design author owns the connected candidate and all its operating/fault cases. |
| B | Astra or another independent checker challenges the assumptions, calculations and complete candidate. It does not author the correction it accepts. |
| C | One clearly scoped P0 supporting task, such as the CAN fault correction or a source/thermal bound, coordinated with the power author and on separate files. |

The three-worker limit includes all active authors and reviewers; the coordinator is additional. There must be one writer for each owned file. Leave a slot unused if no independent P0 task is ready. Do not resume the old allocation automatically.

Keep one authoritative operating envelope and budget. It must connect sources, charging, storage, converters, loads, feed and return conductors, connectors and protection. Use consistent boundaries for voltage, current, losses and heat. Cover required simultaneous operation, startup, docking, charging, all-transmit, relevant temperatures and component tolerances, and the required fault combinations. Do not stack mutually exclusive states or omit permitted combinations.

For every correction, trace its effects through that complete path before calling it a candidate. Recheck changed load, voltage drop, ground current, protection coordination, thermal limits and required service together. A typical value or typical thermal shutdown is not a guaranteed protective limit. Keep model results, printed guarantees and measurements distinct.

Use existing later-layer drafts as inputs. A narrowly necessary circuit edit, component check, fit check, interface correction or composition test may be brought forward solely as a named prerequisite of the current power gate. It must have a stated reason and acceptance check. This is not permission to restart general work in Layers 5–12 or to count those layers as complete.

## 5. Define and enforce the Layer 4 exit gate before redesigning

Use the existing acceptance criteria and make their power implications explicit. Do not weaken them to produce a completion label. Layer 4 cannot be declared complete while an unresolved fact could overturn the selected architecture, its mandatory service, its safe operating envelope or its physical feasibility.

The power portion of the exit gate requires:

- One coherent selected design, with precise circuit/generator changes and compatible interfaces. Separate uncomposed drafts are insufficient.
- Every current desk-fixable power defect corrected and verified against its actual failure case, including the connected consequences of each correction.
- Reproducible calculations tied to the actual candidate and source inputs; explicit margins, uncertainty and applicable operating conditions.
- Independent acceptance of the decision-critical corrected design. Preserve every earlier negative verdict. A coordinator sign-off or an exhausted review allowance does not resolve an outstanding independent blocker.
- No architecture-defining dependency hidden under "conditional", "supplier test", "closed on paper" or a later layer number.
- A stable candidate that passes the applicable existing integration gates on the revision being accepted.

Separate later qualification from unresolved feasibility. A later test may confirm a design already supported by conservative evidence, where the existing layer criteria permit this. If its outcome decides whether the architecture works at all, it is still a current blocker. Identify the specimen, measured quantity, pass limit, required capability and owner; do not claim a planned test has passed.

We have no in-house electronics engineer, and supplier engineering or firmware support has not been secured. Prepare a concrete request when external work is essential. Do not assume NextPCB, Seeed or an unnamed engineer has accepted it. Do not contact anyone or buy hardware without the required authorisation.

## 6. Converge quickly without forcing a pass

- Reproduce each material failing case before changing the design. Prefer the simplest supported correction with useful margin and the fewest new uncertain dependencies. Do not tune a model to match historical numbers.
- When a component's missing guarantee is the obstacle, first make a bounded comparison of practical design alternatives. Select a route within the approved requirements where evidence supports one. Endless searches for the same unavailable limit are not progress.
- Give the independent checker the complete candidate and its assumptions, not a request to confirm the author's conclusion. Use one focused review and a targeted recheck of substantive corrections and their affected interactions.
- If the same failure survives two attempts, stop repeating that method. State the counterexample and change the circuit approach or identify the exact external action needed. A changed design still needs independent checking; do not convert a failed review into acceptance to honour a run budget.
- Generate and bind documentation after the technical inputs stabilise. Use the existing tools and registers; do not create another governance framework. Preserve required evidence without adding cosmetic work to the critical path.
- Freeze one coherent candidate, run affected checks and the required suite, and integrate without concurrent edits to its bound inputs. Reuse valid evidence only where its assumptions and content bindings remain valid. Never relax a test to make the candidate green.

## 7. Restore strict layer order

Layer 4 is the active layer. Layers 5–12 remain paused except for the explicitly bounded prerequisites above. Existing work is retained as provisional evidence, not lost or accepted by implication.

After the full Layer 4 gate passes, proceed to Layer 5; after Layer 5 passes, proceed to Layer 6, then 7, 8, 9, 10, 11 and 12. Keep the repository's firmware/documentation and physical subgates visible. Do not skip a blocked layer merely to keep workers busy. Worker parallelism is within the active layer and its indispensable prerequisites.

For each layer, name its inputs, scope, exit criteria and accepted revision. Check relevant downstream feasibility constraints before accepting an upstream choice. Detailed design can reveal new evidence later: if it invalidates an accepted assumption, reopen the affected gate and pause dependent progression while correcting it. Do not leave upstream acceptance unchanged while patching around a contradiction downstream.

A set number, promoted commit, test count or completed document is not a completed layer. Report "100%" only when that layer's actual scoped acceptance criteria are met. Fabrication release remains a separate gate.

## 8. First checkpoint and reporting

Your first useful checkpoint should be within 30 minutes of execution starting, subject to actual recovery constraints. Report:

1. Which old workers and processes are stopped, where their work is saved, and any exception.
2. The verified baseline and the short P0 blocker list.
3. The author, independent checker and supporting assignment.
4. The first circuit correction/reproduction being worked and the next concrete artifact.
5. The critical path and an evidence-based time range, separating desk execution from external waiting.

Thereafter give a brief checkpoint at least every 45 minutes or at a material result. State defects actually eliminated, new failures discovered, current critical-path work and the next deliverable. Label measured durations and estimates. If a checkpoint slips, identify the cause and change the execution approach where needed; do not simply move the finish time again.

ASAP means prioritising a defensible engineering result and removing avoidable work. Do not promise that every physical unknown can be solved by tonight, and do not trade correctness for a deadline. If desk work reaches a real external blocker, deliver the exact bounded decision or experiment immediately and say the layer remains blocked. Continue other P0 work in the same layer; do not restart downstream work.

Deliver one connected, independently checked power candidate and its honest gate verdict. Then advance layer by layer under these rules.

---

## 16. Review of the P0 execution plan: proceed after four targeted amendments (calibration and layout bounds need a feasibility basis; the integration order and one combined base; preserve work and start engineering beside the clerical work; the external closure path made actionable) (as received)

# MeshSat P0 execution plan — targeted review and amendment

## Decision

**Proceed after the targeted amendments below. Keep the P0 plan; do not start another planning cycle.**

The proposed allocation follows the owner's intent: stop current assignments, preserve their work, give F01 an author, confine three workers to the connected power design, retain independent checking, and pause downstream layers.

The source is still an approval-stage plan. It explicitly says nothing has been stopped yet. This review does not establish that any worker has stopped or any circuit has been corrected.

## Evidence and scope

Reviewed the active plan in `Pasted text(20261005-123653).txt`, lines 11–169, dated 5 October 2026, 14:35 CEST. The superseded appendix is historical context, not an active task queue.

Source SHA-256: `771502d31632d84d60e57b65994f30e80151a7b0c016a9f2563fe68c5de82cff`.

This is a dependency and execution-plan review. I have not independently inspected the named branches, component specifications, calculations, command implementations or V6 report. The numerical margins and proposed circuit alternatives remain unverified here.

## Required amendments

### 1. Calibration and layout targets need a supported feasibility basis

**P1 — verification gap.** P0-1 proposes replacing a detector's missing printed accuracy with per-unit calibration and a Layer 12 test row (lines 60–68). P0-2 similarly proposes plane-resistance bounds, and section 7 carries a layout bound as a condition (lines 69–73, 153–156).

These can be legitimate engineering routes, but writing a calibration procedure or a resistance target does not demonstrate that the design can meet it. Before crediting a correction, establish the calibration uncertainty and applicable operating envelope, and the realizability of the proposed conductor geometry. Account for relevant drift, temperature, tolerances and interconnections in the actual acceptance bound.

If a measurement is needed to decide whether the architecture is feasible, retain the architecture blocker. If conservative evidence already establishes feasibility and a later test merely verifies production implementation, record that narrower qualification obligation. Do not reject calibration as a method; do not treat a future calibration as a completed proof.

**Acceptance:** the author and checker can identify the evidence establishing the claimed bound and which remaining tests confirm implementation rather than decide feasibility.

### 2. Correct the integration order and align the authors' inputs

**P1 — confirmed ordering inconsistency, plus an input-consistency risk.** P0-6 is described as final composition on the frozen candidate (lines 85–86), while Slot A is assigned P0-1, P0-2, P0-6 and then P0-7 (lines 113–115). This places the final composition before the solar-guard work it must include. Slot C also starts from a different branch base (lines 123–128).

Complete the selected solar-guard correction and all other material P0 changes before final composition, independent acceptance and freeze. Perform useful composition checks incrementally, but call only the complete result final. Give both authors the same verified combined baseline, including round 16, or explicitly bring the required selected inputs into each branch before editing them. Keep the shared case definitions under one writer with clear handoffs.

**Acceptance:** the final candidate contains every selected correction, the check evaluates that combined state, and no technical correction is scheduled after its final composition or acceptance.

### 3. Preserve actual work and shorten the administrative critical path

**P2 — checkpoint and scheduling gap.** The recovery step lists tips, statuses and untracked files without explicitly backing up the modified file contents. The serial estimates are 20 minutes for stopping, 25 for the list and 15 for briefs, while the first checkpoint at 30 minutes promises assignments and a reproduction (lines 38–49, 160–166).

Save staged/unstaged diffs and relevant untracked contents, in addition to metadata. Stop the relevant parent/launcher processes as well as their children so they cannot relaunch work. Record the observed state at the time of stopping.

After the safe checkpoint and essential baseline verification, launch the first F01 reproduction and CAN task. The coordinator can finish register formatting alongside that work. Use the 30-minute checkpoint to report what has actually happened; do not wait an hour to start engineering merely to finish administrative text.

**Acceptance:** interrupted work is recoverable, no cancelled assignment is running or scheduled to relaunch, and the first checkpoint distinguishes completed recovery from active engineering and remaining setup.

### 4. Make the external closure path actionable immediately

**P2 — completion dependency.** The plan explicitly expects U-01, U-02 and U-04 to keep Layer 4 blocked even after its estimated 12–16 hours of desk work (lines 94–99, 134–142, 163–167). That is honest, but it is not an ETA for full Layer 4 closure.

At the first checkpoint, state for each claimed architecture blocker: the exact missing fact; why existing evidence does not establish it; the concrete owner decision or specimen/measurement needed; expected cost if known, or how the quote will be obtained; and who must provide the capability. Reuse the existing engineering work. Do not assume a supplier has accepted the job, and do not send requests or make purchases without authorisation.

Include P0-7 in the remaining desk schedule. Keep the estimate for a checked desk candidate separate from the unknown date for full closure. Strict layer order means downstream layers remain paused if an architecture-defining external fact remains unresolved.

## Paste into Claude's plan feedback

```text
Keep this P0 plan and make only these bounded amendments before the normal execution handoff. Do not start another broad planning round.

1. Calibration and layout bounds are proposed means of correction, not evidence by themselves. For P0-1, establish the calibration uncertainty and valid operating envelope before claiming an accuracy bound. For P0-2, demonstrate that the resistance bound is physically realizable with the selected geometry and tolerances. If a measurement decides feasibility, the Layer 4 blocker remains open; a Layer 12 row or layout constraint cannot close it by declaration.

2. Correct Slot A's order: P0-7 and every other selected technical correction must precede final P0-6 composition, independent acceptance and freeze. Both authors must use the same verified combined inputs, including round 16, before editing. Keep one writer for the common operating-case definitions. Early composition checks are useful; only the complete candidate is final.

3. The stop checkpoint must preserve modified file contents and staged/unstaged diffs, not just tips/status lists. Stop launchers as well as children. Once that checkpoint and the essential baseline verification are complete, start F01 and the CAN correction while the coordinator finishes clerical register work. The first checkpoint reports actual progress; it is not a reason to delay engineering for a full hour.

4. At the first checkpoint, make U-01/U-02/U-04 actionable: exact missing fact, existing evidence gap, concrete decision or measurement, required capability, and cost/quote status. Keep correspondence unsent and purchases unauthorised. Include P0-7 in the estimate. State clearly that 12–16 hours estimates a checked desk candidate, not full Layer 4 closure while external architecture blockers remain.

Then execute the approved stop-and-preserve step and the P0 assignments. Preserve the three-worker limit, strict layer order, independent acceptance and the original owner requirements. Do not soften any gate or restart the cancelled queue.
```

---

## 17. Second review of the revised plan: READY to approve for execution; the baseline watchpoint; 14 to 18 h is a desk candidate, not Layer 4's closure (as received)

# MeshSat P0 — revised plan check

## Decision

**READY to approve for execution.** The revised plan addresses the four requested amendments. No further planning round is needed on those points.

This verdict concerns the execution plan. It does not accept the power design, verify the proposed calculations or authorise fabrication, purchases or external messages. Power closure remains blocked as the plan reports.

## Scope

Reviewed the active plan in `Pasted text(20261005-124452).txt`, particularly its revised recovery, correction, assignment and timing sections. The superseded appendix remains historical context.

Source SHA-256: `39fe02a9a439f023529b6877b821e331fc96de3584176f825e3927b9a06dec15`.

Method: compared the revised text with the four amendments in the preceding plan review. No repository operations, hardware calculations, test runs, vendor claims or process states were independently verified here.

## Amendment check

| Requested change | Revised evidence | Result |
|---|---|---|
| Calibration and layout targets need a supported feasibility basis. | Lines 76–92 require calibration uncertainty and operating-envelope evidence, realizable conductor geometry and hot-corner resistance. A measurement that decides feasibility keeps the Layer 4 finding open. | Addressed in the plan; engineering proof still owed. |
| Solar correction must precede final composition, with consistent author inputs. | Lines 104–112 make P0-6 final only after P0-7 and all selected corrections. Lines 132–160 establish a common combined baseline and one writer for shared case definitions. | Addressed in the plan; integration still owed. |
| Preserve actual unfinished work and start engineering alongside clerical work. | Lines 43–60 explicitly preserve staged/unstaged diffs and untracked contents, stop parents/children, check for relaunches, and start F01/CAN work after the checkpoint and essential baseline preparation. | Addressed in the plan; checkpoint and launch evidence still owed. |
| Make external closure dependencies actionable and distinguish desk work from full closure. | Lines 188–205 require missing facts, specimens/limits, capability, owner and cost/quotation status at the first checkpoint. The revised estimate includes P0-7 and labels the result a desk candidate. | Addressed in the plan; decision packets and external evidence still owed. |

## What should happen next

Approve execution through Claude's existing handoff. The first checkpoint, about 30 minutes after approval, should show:

1. Which old assignments are stopped and where their recoverable work is saved.
2. The verified combined baseline and actual status of the F01 and CAN tasks.
3. The next concrete engineering artifact, with any setup delay identified.
4. Actionable U-01, U-02 and U-04 dependencies, with E11-29's qualification obligation kept distinct.

The first checkpoint is an observation of progress, not a promise that every preparation step must already be finished. The plan itself estimates about 40 minutes for stopping, baseline preparation and launch.

One execution watchpoint: if baseline checks fail on a known defect that the P0 authors are assigned to fix, distinguish that from a new merge regression. Preserve the failing result and its owner; do not weaken a test or let the need for an initially green baseline create a circular wait for its own correction. Investigate this only if it actually occurs.

## Timing and remaining limits

The estimate is now **14–18 hours for a connected, independently checked desk candidate**, conditional on the anticipated review outcome. That estimate has not been validated by this review.

Full Layer 4 closure has no supported completion date in the plan: U-01, U-02 and U-04 are still identified as architecture-level external dependencies. Under the owner's strict sequence, Layers 5–12 stay paused while such blockers remain unresolved, except for explicitly named prerequisites of the active gate.

The report says the firmware box jobs finished, but their review remains incomplete. Saving those results preserves work; it does not produce a firmware verdict or justify restarting that cancelled task now.

The next useful evidence is execution and a corrected circuit candidate, rather than another revision of this plan.

---

## 18. Review of P0 checkpoint 1: continue the authors; finish the external decision packet (U-02's per-mode reconciliation and the mock-up's sum, U-04's evidence route apart from the whole-kit release, U-01's two kinds of evidence) (as received)

# MeshSat P0 checkpoint 1 — review

## Decision

**Continue the current P0 authors. No new plan or worker restart is needed.** The checkpoint reports the intended change in allocation: previous work preserved, rented compute stopped, a common power baseline established, and two authors on F01/all-transmit and CAN fault corrections. Astra is correctly shown as queued until there is a selection to assess.

No new power correction is yet reported as independently accepted. Power-design closure and fabrication release remain BLOCKED.

## Evidence and scope

Source: `MESHSAT-P0-CHECKPOINT-1-2026-10-05-1530.md`.

SHA-256: `270de3a1e12283bd057d61dc2b7653497aa7da4b41888856942170385bcbc846`.

I reviewed the checkpoint against the approved execution plan. I did not inspect the remote processes, backups, repository, V6 report, datasheets or test procedures. Process states and test results below are the coordinator's reported evidence, not independently observed execution.
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

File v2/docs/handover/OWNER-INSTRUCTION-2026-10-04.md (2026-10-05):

# The owner's instructions of 4 October 2026: the execution constitution, his reviews of the plans and of the evening's status report, and the continuations

Filed as received (MESHSAT-1357), byte for byte inside each part below, including the owner's own typography. Nothing here is
edited. Part A of the first instruction is the standing execution constitution, extracted as `v2/docs/EXECUTION-CONSTITUTION.md`
(the one authoritative process text; one dash written out there). The live plan that applies them is `v2/docs/EXECUTION-PLAN.md`,
entry of 4 October 2026 14:25 CEST.
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

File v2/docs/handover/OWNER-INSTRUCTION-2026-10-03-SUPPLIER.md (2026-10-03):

# Owner instruction, 3 October 2026: the supplier engineering handover (an amendment to the running plan)

Received in the coordinating session on 3 October 2026, filed as received; it amends the plan of 2 October (`OWNER-INSTRUCTION-2026-10-02.md`) from this point.

## The covering note

Read the attached prompt and apply it as an amendment to the running plan. Preserve current workers, completed calculations and accepted baselines.
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

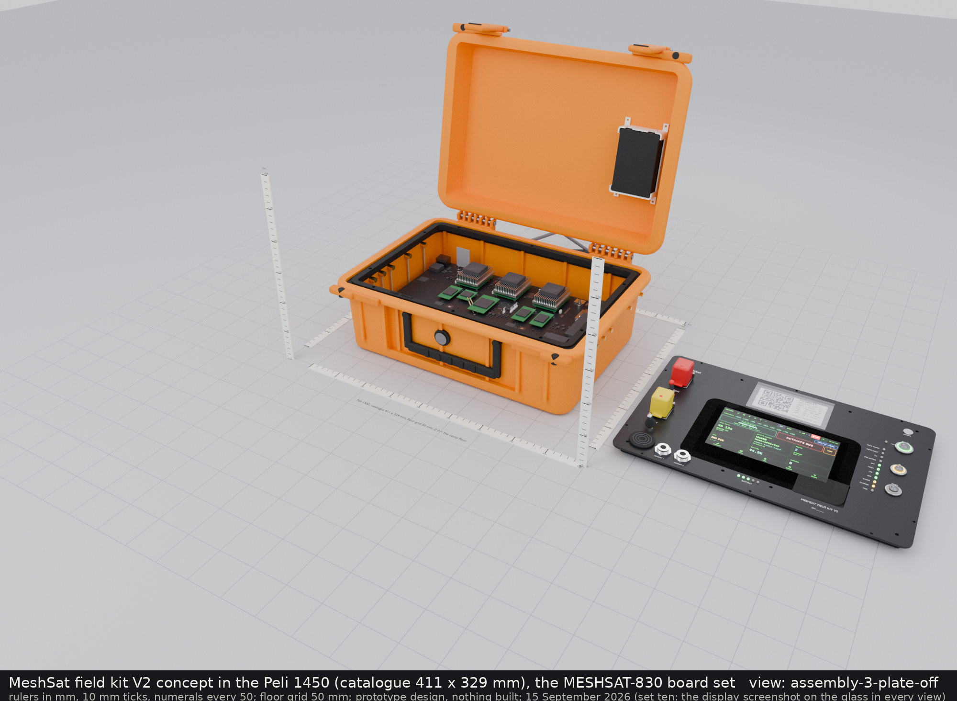
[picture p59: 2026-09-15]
v2/images/concept-1450/set-ten/03-assembly-3-plate-off.png

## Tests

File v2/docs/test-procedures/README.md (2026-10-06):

# Test procedures for the prototype qualification (MESHSAT-1357; the supplier's phase 2)

**Status: PROPOSED, for the supplier to review and agree before execution.** Written 3 October 2026 under MESHSAT-1357 on the
owner's instruction of the same day (`v2/docs/handover/OWNER-INSTRUCTION-2026-10-03-SUPPLIER.md`). The MeshSat field kit V2 is an
**unbuilt prototype design**: no board has been fabricated, assembled, powered or measured, and nothing in these procedures has
been run. They were written by an AI agent session from the project's records; none of them is an electrical engineer's
sign-off, and none has been reviewed by a test laboratory.

**What this folder is.** The records already specify each experiment the power design still needs (what to measure, on which
specimen, against which limit, and what a result may be used for). This folder turns those specifications into procedures a
supplier's engineers can price, review, correct and run. It changes no specification: every pass condition is quoted word for
word from the register row or the record that owns it, and `tp_check.py` holds each quote to its source in this tree. Where a
procedure needs a figure no record states, it writes `TBD (owed by <row>)` naming the register row that owes it; it never
invents the figure. Method details that the records leave open (a sampling rate, the order of runs, a proposed instrument
class) are marked as this folder's **proposal**, for the supplier to accept or replace.

The entry page of the supplier package is `v2/docs/handover/supplier/SUPPLIER-HANDOVER.md`; its sections 5 and 6 explain why
these experiments exist. The route table these procedures implement is section 5d of
`v2/docs/records/l4e9/L4-POWER-ARCHITECTURE.md`; each board A specimen's own block is section 17d of
`v2/docs/records/l4e11/L4E11-SOURCE-ONLY-AND-ENTRY.md`; the acceptance of every row is in
`v2/docs/records/l4e9/DOWNSTREAM-REGISTER.md`.

## 1. The procedures

| Procedure | File | Register rows | What it decides | Performer (from 5d) |
|---|---|---|---|---|
| TP-TH1 | `v2/docs/records/l4e12/T-H1-PROCEDURE-DRAFT.md` (written earlier, not in this folder, not rewritten here) | R-104, R-151 | U-02: the sealed case's conductance per required mode | an engineer, on a bench |
| TP-E11-29 | TP-E11-29.md | R-159 | D-14's installed thermal path and junction limit of the three battery FETs Q39, Q40 and Q42 (its acceptance awaits a correction and the supplier's agreement: its section 8; not to be run yet) | an engineer, on a bench (the body diode's VSD method) |
| TP-E11-30 | TP-E11-30.md | R-160 | D-14's docking pulse: the whole hot waveform in one body diode | an engineer, on a bench (a capacitor-discharge rig) |
| TP-E11-36 | TP-E11-36.md | R-182 | D-14's RDS(on) allowance at VGS -8.5 V and a 150 C junction | an engineer, on a bench (an oven to 150 C, a pulsed Kelvin reading) |
| TP-E11-37 | TP-E11-37.md | R-183 | BATDRV with the three battery FETs on one gate node, their current sharing and junctions: the three (S1), or the pair at its fallback or one FET with a case heat path (S2) | an engineer, on a bench |
| TP-E11-31 | TP-E11-31.md | R-161 | U-04: source-only start and the held states on the BQ25730 | an engineer, on a bench |
| TP-E11-38 | TP-E11-38.md | R-184 | D-15: the eFuse U42 and the dock's VSYS branch through cases (a) to (h) | an engineer, on a bench |
| TP-E11-35 | TP-E11-35.md | R-179, R-188 | the mixer fans' start current and PWM level, and the firmware's stagger (E11-35, E11-39) | an engineer, on a bench |
| TP-SOLAR | TP-SOLAR.md | R-176, R-189, R-174 | D-10, D-11 and D-16: the solar input guard's thresholds and waveforms at U5's pins, and the sense in operation | an engineer, on a bench; CS116 and CS115 a MIL-STD-461 laboratory |
| TP-EPAPER | TP-EPAPER.md | R-185 | U-02's missing storage qualification of the e-paper (M6, M7) | an engineer with an oven, or a laboratory |
| TP-CELL | TP-CELL.md | R-168, R-169 | U-01's Saft route: the one-cell limited sample qualification | a laboratory |

**One warning carried by TP-SOLAR.** The drafted solar guard is known, on the desk model, to FAIL its own row at a fault at the
connector: U5's sense pins reach past their absolute maximum (handover row P1, task P1-1). TP-SOLAR therefore measures the
supplier's **corrected** network (the output of phase 1's task P1-1), and says how to treat the drafted one if it is ever
stepped.

**Rows of 5d's route table not written here**, each with its reason (machine-read by `tp_check.py`, which requires every 5d row
to be covered exactly once):

<!-- tp-index
external: TP-TH1 | v2/docs/records/l4e12/T-H1-PROCEDURE-DRAFT.md | R-104, R-151 | T-H1 (R-104, R-151; T-H1-PROCEDURE-DRAFT.md)
not-covered: The HL18650V lot soak (R-103, R-47; route (II) only) | the HL18650V route (II) is an alternative only; its soak is specified in 5d and L4-E10 15e and is not part of this set's request
not-covered: The fit mock-up (R-167) | a printed geometry check owned by Layer 7, no instrument and no pass line beyond the fit itself
not-covered: The documentary alternatives (the makers' statements) | not an experiment: the owner sends the drafted requests; a maker's printed limit closes a row for every lot
-->

- **TP-TH1** is the existing draft `v2/docs/records/l4e12/T-H1-PROCEDURE-DRAFT.md`; it is the model the others follow for depth.
- **The HL18650V lot soak** (route (II) only) is not written: it serves an alternative cell, not the selected route.
- **The fit mock-up** (R-167) is a print in the pocket, Layer 7's.
- **The documentary alternatives** are the makers' statements; a returned maker's limit closes its row for every lot and makes
  the matching procedure here unnecessary for that row.

## 2. How each procedure is laid out

Every TP file has the same eleven sections: (1) purpose and the decision it settles, with its register row; (2) the specimen and
what transfers, quoted from 5d and 17d; (3) safety; (4) equipment, with the accuracy each measurement needs and how that accuracy
follows from the pass limit and the uncertainty budget (an instrument class is named, never a brand); (5) setup and measurement
points; (6) the steps; (7) the data to record, as a table template; (8) pass, fail and inconclusive, quoted from the register or
the record; (9) the uncertainty budget's terms; (10) the consequence of a fail and the re-test triggers; (11) the authorisation
and purchases needed, quoted from 5d (nothing has been bought).

A metadata block at the top of each file (an HTML comment) names its id, title, register rows, L4-E11 rows and 5d route rows for
the checker. A quote sits between an opening HTML comment marker ("q", naming its source and, for a table cell, its row and column)
and a closing one ("/q"); the checker compares it with the source cell or text. A quote is the record's wording, including its own cross-references (section numbers such as "16b" or "17d"
are sections of the quoted record).

## 3. The verdict rule shared by every procedure

The records state the rule for a reading against a limit in two places:

<!-- q src="v2/docs/records/l4e11/L4E11-SOURCE-ONLY-AND-ENTRY.md" -->
> **Measurement uncertainty:** the K-factor within 2 %, the heating power within 1 %, the air within 1 K, stated as an expanded
> uncertainty on Zself + 2 Zmut; a reading passes when it plus its ACHIEVED expanded uncertainty is under the limits of E11-29
> (round 14, V2R-m4: the supplier's achieved U, not a fixed figure).
<!-- /q -->

<!-- q src="v2/docs/records/l4e12/T-H1-PROCEDURE-DRAFT.md" -->
> Per point: **pass** when the reading less its expanded uncertainty is at or over the line's need (the reading at or over the
> threshold below); **fail** when it is under; **inconclusive** when the endpoint is not met
<!-- /q -->

So, in every procedure here (the general form of those two sentences; nothing in it lowers a limit):

| Result | Against an upper limit L ("at most", "under") | Against a lower limit L ("at least", "over") |
|---|---|---|
| **PASS** | the reading plus its expanded uncertainty U is at or under L ("at most") or under L ("under") | the reading less U is at or over L ("at least") or over L ("over") |
| **FAIL** | otherwise, on a valid measurement. A reading that is itself inside L but whose band reaches past it does not pass: it is reported as FAIL, marked "within uncertainty", as T-H1 section 6 treats it; a repeat at a smaller U is a new run, and the first run stays in the record | the same |
| **INCONCLUSIVE** | a validity condition of the procedure is not met (the specimen differs from its block, the operating point is not held, an instrument is out of calibration or its uncertainty is not achieved, the endpoint is not reached); the run is repeated; an INCONCLUSIVE run is never a pass | the same |
| **RECORDED** | the record asks for a value and states no limit: the value and its U are filed and no verdict is given | the same |

- **U** is the expanded uncertainty at a coverage factor k = 2, as T-H1 uses it, combined from the standard uncertainties of the
  budget's terms by root-sum-square where they are independent (the method of the ISO Guide to the Expression of Uncertainty in
  Measurement, JCGM 100:2008; not held in this tree). Each procedure lists its terms in its section 9.
- **A planning target, this folder's proposal:** an instrument chain whose U is at most a quarter of the margin it judges (a
  test uncertainty ratio of 4:1, the usual calibration-laboratory practice). It is not a validity condition: a larger U only makes
  a PASS harder to reach. Where a record states an accuracy (the 17d blocks do), the record's figure governs.
- **Every instrument** carries a calibration traceable to national standards and inside its interval; its model class, serial
  number and calibration date are recorded with the run.

## 4. What a result is, and what it is not

<!-- q src="v2/docs/records/l4e9/L4-POWER-ARCHITECTURE.md" -->
> **The rule.** An evidence build proceeds under its own scope; the design and production release stays held until the
> measurements pass; a row is not closed because it has an owner and a future test. A sample result is evidence for that lot and
> that sample, never a production limit; only a maker's printed limit closes a row for every lot. Purchases and outside contact
> are the owner's: nothing here is bought or sent.
<!-- /q -->

<!-- q src="v2/docs/records/l4e11/L4E11-SOURCE-ONLY-AND-ENTRY.md" -->
> So **a coupon's thermal result transfers only where the final board's thermal boundaries are shown no worse by a named rule, and
> a sample's pulse result is prototype evidence for that lot and those conditions, never a production limit or an extension of the
> maker's guarantee.**
<!-- /q -->

## 5. Authorisation, acceptance and the record to keep

- **Authorisation to perform** a procedure (the bench, the people, the spend on parts and fixtures) is the owner's, as each 5d
  row states in its Authorisation column. Nothing here has been bought, sent or run.
- **Acceptance of a result** goes through the coordinator's check of the filed record against the register row and the record
  the procedure quotes, as T-H1 section 0 sets out for its own points. The owner's authorisation does not accept a result, and a
  passing result authorises nothing further.
- **No limit is relaxed to make a run pass.** A run that fails is reported as failing, with the consequence its section 10
  quotes.
- **The record to keep**, for every run: the raw instrument files; the specimen's identity (part numbers, lots, reels, date
  codes, the coupon's fabricator, stack-up and copper weight); photographs of the specimen and of every measurement point; the
  instruments' classes, serial numbers and calibration dates; the ambient and chamber logs; the reduction (a script or a
  worksheet) and its output; the verdict per pass line with the reading, its U and the limit; who ran it, where and when, under
  which authorisation. The filled table templates of each procedure's section 7 are the summary, not a replacement for the raw
  files.

## 6. Safety that applies to every procedure

Each procedure's section 3 names its own hazards. Common to all: the laboratory's own electrical-safety rules and permits apply
and take precedence over anything here; supplies are current-limited to the run's need; a specimen is never left energised
unattended unless the procedure provides an automatic abort; chambers and ovens are used within their ratings, with burn
protection for parts handled hot; a lithium-ion cell or pack is handled under the laboratory's battery-safety rules (a fire-rated
enclosure, voltage and temperature monitoring with automatic cut-off, an exhaust for venting gases). No procedure here is to be
run on the owner's kit hardware or by the owner.

## 7. The bring-up page

`v2/docs/PCB-BRING-UP.md` carries, since 3 October 2026, the supplier's bring-up procedure for the first prototype of each board (A,
B, C, D, E, E5 and P): per board the drafts the prototype is built with (each with its register row, and what may not be powered
when a known-defect correction is missing), the first power-up on current-limited supplies, the rails and their bands, the checks
before the next board is connected, the firmware and register writes, the hand-offs to the procedures of this folder and to the
register's bench rows, and the stop conditions. It describes the design with the drafts applied, which is not the committed
schematic, and is marked PROPOSED like every procedure here.

The page was generated whole by `tools/rules_render.py` (rule TST-001 compares it with the boards' intent files). The procedure is
written by hand ABOVE the renderer's marker, and the renderer keeps that part unchanged at every render (`_with_bringup_preface`);
only the rail inventory under the marker is generated, so `--check` and TST-001 still judge that part. A page without the marker
renders exactly as before. The page's inputs from branches not in this tree's history (Layer 8's records l8gnd and l8r2, Layer 5's
second round) are copied byte for byte into `inputs/`, each with its branch, commit, source path and sha256 in
`inputs/SOURCES.txt`; the page quotes the copies.

## 8. The checker

`tp_check.py` (run from the repository root: `python3 v2/docs/test-procedures/tp_check.py`) checks every procedure against its
sources and prints the index, the coverage of 5d's route table and every TBD by the row that owes it. It also checks the bring-up
page's procedure (the marker and the generated block under it, the PROPOSED mark and the drafts statement, every quote, path and
TBD, the seven subsections of each board, every register row its tables name) and the inputs' sha256 against `inputs/SOURCES.txt`. Its output is committed as
`tp_check.out` and is regenerated only through the project's `regen_out.py`, which refuses a failed or non-deterministic run.
The test `v2/ecad/tools/tests/test_test_procedures.py` holds the same properties (every procedure names its register row and
the row exists; every pass condition is quoted from its source; every procedure carries the PROPOSED mark; no long dash) and
checks that the committed output is what the script prints. The quotes are checked against the records as they stand in this
tree: if a record's acceptance changes, the check fails and the procedure is re-read before its output is regenerated.

**What a passing check shows, and what it does not.** A passing quote check (`tp_check.py` printing ALL PASS) shows that the
quoted texts match their sources; it does not approve any procedure to run. Every procedure stays PROPOSED until the supplier
agrees it.

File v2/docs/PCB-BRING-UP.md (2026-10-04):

<!-- HAND-WRITTEN above the marker below (MESHSAT-1357, 3 October 2026; checked by v2/docs/test-procedures/tp_check.py). The rail
     inventory under the marker is GENERATED by tools/rules_render.py from each board's intent file and is compared by --check
     and rule TST-001; this part is carried through every render unchanged. -->

# Bring-up of the first prototypes, board by board

<!-- tp-bringup
boards: A, B, C, D, E, E5, P
-->

**Status: PROPOSED, for the supplier to review and agree before execution.** Written 3 October 2026 under MESHSAT-1357 for the
supplier's engineers who build and bring up the first prototypes (the supplier package, phase 2). Prototype design: **no board has
been fabricated, assembled or powered**, and nothing here has been run. Written by an AI agent session from the project's records;
it is not an electrical engineer's sign-off.

**This page describes the design WITH the drafts applied, which is not the committed schematic.** The generators and netlists
committed in this tree are the boards before the Layer 4 and Layer 8 drafts: every draft named below is a release-guarded apply
script that no generator carries yet. A first prototype is built from the regenerated boards once the drafts it needs are
released and applied; each board's section 1 states which drafts the prototype must carry, and what may not be powered when one of
them is missing. Appendix A (under the marker at the end) is the rail inventory as the committed intent files declared it at the
last render, before any draft; where a draft adds or changes a rail, this page names it with its figure from the draft's record.

**Sources.** The Layer 4 records in this tree (`v2/docs/records/l4e9/L4-POWER-ARCHITECTURE.md` section 3, the change list in
application order; `v2/docs/records/l4e9/DOWNSTREAM-REGISTER.md`, every row's acceptance; `v2/docs/records/l4e11/L4E11-SOURCE-ONLY-AND-ENTRY.md`),
`v2/docs/ARCHITECTURE.md` section 4.3, and four inputs from branches not in this tree's history, copied byte for byte with their
sha256 and source in `v2/docs/test-procedures/inputs/SOURCES.txt`: Layer 8's records l8gnd (`fnd/l8gnd` at 226e9143) and l8r2
(`fnd/l8r2` at a441651a), and Layer 5's second round (`fnd/l5r2` at 6902db8f: `pcb_interfaces.yaml`, `HW-FW-CONTRACT.md` and its
record). A figure no record states is marked to be determined, naming the register row that owes it. Method details the records leave open are marked as this page's
proposal.

## 0. The order the boards come up, and the rules for every step

**The order** (proposal; each step only after the previous one has passed its stop conditions):

1. **E5**, the dock block: no power; continuity, isolation and contact resistance (section E5).
2. **P**, the pack board, on a cell simulator, never on cells first (section P).
3. **C**, the panel board, alone on a bench 5 V supply, with its controller's firmware loaded (section C).
4. **A**, the power board, alone on bench supplies (section A).
5. **D** on A over the mezzanine harness and the 5 V lead (section D).
6. **B** on A over the rail leads and the A to B ribbon, then **C** on B over the panel ribbon and to A over the MAIN lead (sections B
   and C).
7. **E** alone on bench supplies, then E with A through E5 (section E).
8. The pack (P with its cells) on E's J_BATT, the stack seated on E5, only after the docking pulse has been qualified (section P).

**Rules for every step.**

- **Current-limited supplies, in two stages.** Stage 1: the limit set just above the expected no-load current with every switched
  load at its power-up state (`v2/docs/ARCHITECTURE.md` 4.3's line-state table, quoted in section A). The records do not itemize the
  power path's quiescent draws, so the expected stage-1 current of each board is owed by the budgets row, R-51 (the record's own
  statement is quoted below); stage 1 records it as the board's baseline. Stage 2: the limit raised to the rail's declared typical
  current (Appendix A's "current limit" column) only for a step that enables a load. A supply that reaches its limit is a short
  until proved otherwise.
- **A derived rail is never applied from the bench**: it is measured where it is made, against its expected value and tolerance
  (Appendix A: plus or minus 5 % of the declared voltage, or the record's tighter band where this page names one).
- **Thermal watch:** every board is scanned with a thermal camera at each stage; a part that heats with no load to explain it is a
  stop. Temperatures are recorded, not judged here (the thermal acceptance belongs to T-H1 and the TEST-PLAN rows).
- **Every stop** leaves the board unpowered and is recorded with the readings that caused it; the step is not repeated until the
  cause is found.

<!-- q src="v2/docs/records/l4e9/L4-POWER-ARCHITECTURE.md" -->
> **The quiescent draws** of the power path are not itemized part by part in any record: the profile carries them inside the
> declared board rows (board A's logic and board E's controller and sensors), the solar stage's own drive and quiescent power
> comes from the panel (M6), and the outlet converter idles only while it is enabled (M2). An itemized list would move the profile
> by the parts' printed quiescent currents; it is not counted here as done.
<!-- /q -->

**The firmware the bring-up needs.** The kit's boot order is the panel controller's (board C's RP2040, FW-C01); during a board's
bring-up alone, a bench I2C host on the kit bus performs the same writes in the same order. The contract rows, from Layer 5's copy:

<!-- q src="v2/docs/test-procedures/inputs/l5r2-HW-FW-CONTRACT-6902db8f.md" row="FW-C01" col="Firmware obligation" -->
> 1. PI_KILL low; 2. PI_SHDN_REQ released; 3. read ZEROIZE_SW and the wipe-pending record, complete any pending wipe; 4. every
> expander's outputs before its configuration (FW-A08); 5. the charger (FW-A01 to A03, A16, A17, A18); 6. SLOT_EN1..3 one at a
> time, each after the keeper's held level has been read and adopted (FW-C02; with the hold applied, record l8gnd). Never the
> RP2040-E5 USB fix; a BOOTSEL activity mask of 0 or GPIO25 only
<!-- /q -->

<!-- q src="v2/docs/test-procedures/inputs/l5r2-HW-FW-CONTRACT-6902db8f.md" row="FW-A08" col="Firmware obligation" -->
> Write the OUTPUT registers before the CONFIGURATION registers on every boot; never write DEV_EN (`A:U27.11`, R42 100 k to +3V3,
> ON at power-up) = 0 except as the last act of a shutdown
<!-- /q -->

## Board A

### A1. Preconditions

The prototype carries board A's drafts in the application order of L4-E9 section 3, followed by Layer 8's. Record l8r2 proved the
whole order composes:

<!-- q src="v2/docs/test-procedures/inputs/l8r2-L8R2-KNOWN-DEFECTS-a441651a.md" -->
> L4-POWER-ARCHITECTURE.md section 3's order runs r12, guard, charger (3a), r11 (3b), bank (3c), r138 (3d), u17 (3e). Then come
> l8gnd's gnd002 and hotr1 (3g), this record's d8v3 and vbus20ov, and d8dec31's mainpb last (3h): **OK at every step**.
<!-- /q -->

| Draft (apply script) | Register row | What the prototype carries | If the prototype is built without it |
|---|---|---|---|
| `apply_gen_sch_a_r12.py` | R-01 | R12 12 mOhm and C147 on the front end U2 | R-64's bench line is not judged on that board |
| none: a missing draft | R-03 | the ILIM_HIZ network (H3) to the corrected knee | the firmware's input limit is the derated 4.00 A (R-25, quoted below); R-74 and R-77 are not judged |
| `apply_gen_sch_a_guard.py` | R-124 | U34's restart guard with R14 76.8k | U34 as drawn (its fall up to 8.309 V, Layer 5's `power_line_states`); R-77's guard line is not judged |
| `apply_gen_sch_a_charger.py` | R-157, R-181, R-209 | the BQ25730 with the three battery FETs Q39, Q40 and Q42 (BATDRV; Q42 added by L4-E11's round 9) and the eFuse U42 on J_DOCK pin 1 (VSYS_DOCK) | the drawn BQ25731 with no battery FET and pin 1 on GND: none of TP-E11-29, TP-E11-31, TP-E11-37, TP-E11-38 has a specimen on that board, and board E's auxiliary domain is not fed over the dock (section E) |
| `apply_gen_sch_a_r11.py` | R-04 | R11 8 mOhm | R-60 and R-62 are not judged |
| `apply_gen_sch_a_bank.py` | R-07 | the six 45 mOhm ballasts and Cc2 | R-66 and R-68 are not judged |
| `apply_gen_sch_a_r138.py` | R-05 | R138 5 mOhm | R-79 is not judged |
| `apply_gen_sch_a_u17.py` | R-06 | U17 off the 54 V rail on R227 (POE_VIN) | R-84 is not judged |
| record l8gnd's `apply_gen_sch_a_gnd002.py` | R-191 | the CHASSIS net, its 0 Ohm link R229 to GND and the strap pad H1 | no chassis bond: the bond-resistance reading of section A6 is skipped |
| record l8gnd's `apply_gen_sch_a_hotr1.py` | R-192 | the SLOT_EN keepers U43 with R230 to R232 and C240 | a panel reset drops every slot (V-C02's extended row is not run) |
| record l8r2's `apply_gen_sch_a_d8v3.py` | none in this tree's register (Layer 5's finding L5R2-F05) | the eFuse U44 on board D's 3.3 V (+3V3_D8 on J_MEZZ1 pin 13) | board D's 3.3 V has no branch limiter: board D is joined to A only after its own bench bring-up (section D) |
| record l8r2's `apply_gen_sch_a_vbus20ov.py` | R-48 | **the correction of a known defect** (S-111, supplier task P1-3): VBUS20's over-voltage cut-off, Q41 in series at the VIN_RAW entry (J_VR1 to J_VR4 on VIN_RAW_IN) and U45 | **must not be powered with VIN_RAW over 24 V**, and no fault of section A6 is injected (this page's reading of l8r2 item 2: with Q2 shorted VBUS20 follows VIN_RAW less Q5's body diode, and the cut it would add sits at 24.25 to 25.31 V, under U3's recommended 26 V) |
| d8dec31's `apply_gen_sch_a_mainpb.py` | R-193 (with R-194) | the network at the LTC2954's PB pin, last in board A's round (R248 and C247 after l8r2's drafts, its finding F2-02) | the MAIN press is read through the drawn PB pin |

The firmware input limit on a board without the H3 line:

<!-- q src="v2/docs/records/l4e9/DOWNSTREAM-REGISTER.md" row="R-25" col="Item" -->
> Firmware: IIN_HOST 4.70 A (code 94, 0x5E00, RSNS_RAC 0b), rewritten after every adapter removal; on the drawn board the derated
> 4.00 A
<!-- /q -->

### A2. First power-up

1. **No pack, no other board.** Every board-to-board connector open; J_MAINSW to a bench pushbutton (IF-AC-MAINSW's MAIN lead); a
   bench I2C host on the kit bus at J_AB1 (the pin map is IF-AB-RIBBON's).
2. **VIN_RAW_IN** at J_VR1 to J_VR4 from a bench supply at 12.0 V (Appendix A's VIN_RAW row), stage 1. Expected before MAIN: the
   front end U2 runs once U34 releases, VBUS20 rises, the charger U3 starts, VSYS (the net VBAT) rises; the LTC2954 holds RAIL_EN low,
   so board A's +3V3 stays off. The stage-1 current is TBD (owed by R-51): board A's quiescent draw with every switched load off,
   which no record itemizes.
3. **The charger's first writes** (section A5), then VSYS read against its no-pack line.
4. **MAIN pressed**: +3V3 rises, the expanders U27 and U28 leave reset as inputs, DEV_EN is on by its pull-up, so +5V_DEV starts by
   design; every other enable stays off. Record the input current again.
5. **The pack node from a bench supply, never from a pack:** CELL+ at J_CP1 (and the precharge pin J_PRE1) from a current-limited
   supply at 14.4 V (Appendix A), stage 1. A pack, or any stiff source, on CELL+ produces the docking pulse through one battery FET's
   body diode (242.9 A peak, 33.8 us), which is qualified only by TP-E11-30.
6. **Stage 2, one switched load at a time** through the expanders (section A5's order): each output's enable, its rail measured, its
   current recorded, then off before the next.

The startup the records describe for (B1):

<!-- q src="v2/docs/records/l4e9/L4-POWER-ARCHITECTURE.md" row="power-on under (B1)" col="The figure" -->
> the strap 75.14 % of VDDA; the whole 242.9 A pulse in one FET, TJ 123.3 C from the +70 C air on the stated VF bound, CONDITIONAL
> on VF and ISM hot (E11-30)
<!-- /q -->

<!-- q src="v2/docs/records/l4e9/L4-POWER-ARCHITECTURE.md" row="a source-only start under (B1) (no pack, or both FETs open)" col="The figure" -->
> on held evidence the start ends in VSYS_MIN or in a latch within 3.062 s (the hiccup's 500 ms off and 10 ms retries; the 7th
> failure inside 90 s latches; a re-plug clears it); whether the first window succeeds is not bounded: 0.5 A is an input ceiling,
> not a delivered current (the earlier 502.3 ms withdrawn); E11-31 at -20, 25 and 62.1 C
<!-- /q -->

### A3. Rails

Appendix A's board A table gives every rail the committed intent declares, in dependency order, with plus or minus 5 %. The
records' tighter bands and the drafted rails:

| Rail | Expected | Source of the figure |
|---|---|---|
| VIN_RAW_IN (drafted, J_VR1 to J_VR4) | the bench supply's voltage | record l8r2 item 2 |
| VIN_RAW (behind Q41) | VIN_RAW_IN less at most 28 mV at 5.983 A (Q41 at most 4.6 mOhm) | record l8r2 finding F2-04 |
| VBUS20 | 19.08 to 20.96 V | L4-E9 1a, the FE row (quoted below) |
| VBAT (VSYS), no pack, after EN_OOA 0 | at least 12.054 V | R-161 (TP-E11-31) |
| VBAT (VSYS), charge inhibited, pack node from the supply | VSRN + 150 mV within 2 % above SRN 12.546 V; at least 12.054 V below SRN 12.054 V; at least 11.96 V between | R-161 (TP-E11-31) |
| VSYS_DOCK (drafted, J_DOCK pin 1, behind U42) | VSYS, ramped in 3.99 to 8.75 ms (C237 22 nF) | Layer 5's `power_line_states` VSYS_DOCK |
| +3V3 | 3.30 V plus or minus 5 % | Appendix A |
| +3V3_D8 (drafted, behind U44, J_MEZZ1 pin 13) | +3V3 less at most 14.3 mV at board D's peak | record l8r2 3b |
| +5V_D8 | 4.872 to 5.133 V | Layer 5's R2-16, from board A's intent (stream s99a) |
| CHASSIS (drafted) | joined to GND by R229 alone | record l8gnd 2e |
| SLOT_EN1..3 (drafted keepers) | low at power-up; held high at least 2.547 V, held low at most 0.266 V | record l8gnd 3b |

<!-- q src="v2/docs/records/l4e9/L4-POWER-ARCHITECTURE.md" row="FE" col="Settings and limits (as read; drafted parts named)" -->
> R11 8 mOhm, R12 12 mOhm (drafted); U34 guard R14 76.8k (drafted); VBUS20 19.08 to 20.96 V; efficiency 0.93 declared (C-8)
<!-- /q -->

<!-- q src="v2/docs/records/l4e9/L4-POWER-ARCHITECTURE.md" row="VBAT" col="Settings and limits (as read; drafted parts named)" -->
> 9.688 to 17.375 V (B1); D1 SMCJ18A clamp; no pack: at least 12.054 V;; inhibited: piecewise (15d); Q39, Q40 BUK6Y10-30P; to
> CH_BATQ (drafted;; 0.0934 W at the profile); U42 eFuse to the dock's pin 1,; 1.4713 to 1.8018 A (drafted)
<!-- /q -->

The line states until the panel firmware writes the expanders:

<!-- q src="v2/docs/ARCHITECTURE.md" -->
> | State | Lines |
> |---|---|
> | deasserted, guaranteed | SLOT_EN1..3 (100 k down on A: R30, R34, R38, and the RP2040 pad's reset pull-down); PA_SW_EN, HF_SW_EN, MON_EN, HEAT_EN, D8_EN, POE_SW_EN, PD_SW_EN (4.7 k down, `gen_sch_a.py:1105-1112`, `:1125`, `:1009`: 0.49 V at the expander's 100 uA worst case, under every OFF threshold); POE_EN and PD_EN also need OUTLET_OK; on B: LIME_SW_EN, RB_SW_EN, LORA_ON, ZB_ON, CAM_EN, KSZ_RST, 5G_OFF, 5G_RESET (4.7 k down, `gen_sch_b.py:957`, `:981`, `:1011`) |
> | ON, by design | DEV_EN (R42 100 k to +3V3, `gen_sch_a.py:887`); CHG_INHIBIT low (R21 4.7 k, `:763`), so the charger is not inhibited |
> | radios dark by design | the CM5 on-module radios: U6's off-requests pull up through 10 k into the KILL gates (`gen_sch_b.py:719-741`), so the radios stay disabled until the panel firmware writes U6, and are released (fail open) only if +3V3_DEV is lost while a slot runs (EMCON L3) |
<!-- /q -->

### A4. Before the next board

- **To D** (IF-AD-HARNESS): J_MEZZ1 pin 13 on +3V3_D8 behind U44 (drafted) and its current limit shown (section A6); +5V_D8 inside its
  band at J_MEZZ_PWR1 with D8_EN on.
- **To B** (IF-AB-POWER, IF-AB-RIBBON): each slot rail +5V_S1 to +5V_S3 off with SLOT_EN low, then each in turn at 5.10 V on its own
  enable; +5V_DEV at 5.00 V; +54V_POE off (POE_EN low at power-up); the ribbon's SLOT_EN lines at 0 V before the panel runs.
- **To C** (IF-AC-MAINSW): the MAIN lead's open-circuit level and threshold (Layer 5's R2-18, quoted in section C4).
- **To E through E5** (IF-AE-DOCK): pins 2 to 7 and 11 on GND; pin 1 VSYS_DOCK behind U42 (drafted); pin 8 SHORE_INHIBIT low; pin 12
  DOCK_SPARE held high by R216 (HOT-R1's lost-detector state); VIN_RAW_IN on J_VR1 to J_VR4.
- **The chassis bond** (drafted): R229 the only part between CHASSIS and GND, read four-wire (section A6).

### A5. Firmware and register writes

The charger under (B1), at every charger power-on reset, before any other write:

<!-- q src="v2/docs/test-procedures/inputs/l5r2-HW-FW-CONTRACT-6902db8f.md" row="FW-A23" col="Firmware obligation" -->
> At every charger POR: EN_OOA written 0 first (the printed VSYS accuracy holds only after that write, E11-31); ChargeCurrent
> written for any charge (0 A at POR and after the watchdog's 175 s, so the watchdog is serviced or WDTMR_ADJ set 00); VSYS_MIN,
> EN_LDO, EN_PORT_CTRL, BATFET_ENZ and BATFETOFF_HIZ never written from their power-on values; the device ID D5h checked before
> any write; R-a's bit following the hold flag in every state (S4's exception withdrawn, FW-A19); R-b' under VSYS_MIN (FW-A20);
> IIN_HOST 4.70 A and VINDPM as FW-A16; every ChargeOption write read-modify-write (FW-A17's rule, with the BQ25730's own register
> map)
<!-- /q -->

- On the drawn charger (no (B1)): RSNS_RAC = 0b first (FW-A01), then the input limit (FW-A16).
- IIN_HOST: 4.70 A only on a board with the H3 line; on a board without it the derated 4.00 A (R-25, quoted in section A1).
- The expanders: output registers before configuration, DEV_EN never written 0 except as the last act of a shutdown (FW-A08,
  quoted in section 0).
- The keepers (drafted): before the panel's GPIO13 to 15 are made outputs, each line read and driven at the level read (FW-C02 with
  the hold applied, record l8gnd 3f).

### A6. Hand-off to the test procedures and the bench rows

| Measurement | Procedure or register row | Register row |
|---|---|---|
| the three battery FETs' thermal path and junction limit, if board A's first prototype is the specimen (its acceptance awaits a correction and the supplier's agreement; not to be run yet) | `v2/docs/test-procedures/TP-E11-29.md` | R-159 |
| BATDRV with the three battery FETs, their current sharing and junctions, on the first prototype | `v2/docs/test-procedures/TP-E11-37.md` | R-183 |
| the three modes, the held pack current, the start and D2 | `v2/docs/test-procedures/TP-E11-31.md` | R-161 |
| the dock's VSYS branch through cases (a) to (h), with board E | `v2/docs/test-procedures/TP-E11-38.md` | R-184 |
| the first docking with a pack: the waveform measured and compared value by value with TP-E11-30's tested envelope | `v2/docs/test-procedures/TP-E11-30.md` (its block's comparison rule) | R-160 |
| the front end, the knee, the bank, the outlet, U17's shunt, VBAT's peak at a charge-FET opening | the register's bench rows | R-60, R-61, R-62, R-63, R-64, R-65, R-66, R-67, R-68, R-71, R-73, R-74, R-75, R-77, R-78, R-79, R-84, R-86 |
| the dead-pack and no-pack start | the register's bench row | R-85 |
| VBUS20's over-voltage cut (drafted) | record l8r2's bench rows (quoted below) | R-48 |
| board D's 3.3 V branch limit (drafted) | record l8r2 3b's bench row (quoted below) | none (L5R2-F05) |
| the keepers' power-up and hold | record l8gnd 3h (quoted below) | R-192 |
| the chassis bond | R229 read four-wire, the only path between CHASSIS and GND | R-191 |

<!-- q src="v2/docs/test-procedures/inputs/l8r2-L8R2-KNOWN-DEFECTS-a441651a.md" -->
> **Bench row (Layer 9):** - VBUS20 driven through R241 at its divider: the cut between 24.25 and 25.31 V, the release between
> 23.00 and 23.84 V; - Q2's fault simulated by a link across Q2 with a current-limited 36 V source: the bus at or under 26.0 V; -
> FB's open simulated by lifting R6, with U2 running: the bus at or under 26.5 V and U3's VBUS at or under 26.5 V.
<!-- /q -->

<!-- q src="v2/docs/test-procedures/inputs/l8r2-L8R2-KNOWN-DEFECTS-a441651a.md" -->
> **Acceptance.** J_MEZZ1 pin 13 on +3V3_D8 behind U44 (D8V3: NOT DRAWN today). Bench: board D's 3.3 V shorted at the harness,
> with the current inside 0.224 to 0.269 A and board A's +3V3 held.
<!-- /q -->

<!-- q src="v2/docs/test-procedures/inputs/l8gnd-L8-GND002-SLOTEN-226e9143.md" -->
> **V-C02 extended:** "watchdog reset, RUN reset and SWD reset with three slots running, and the panel's firmware reloaded by SWD:
> no slot rail drops; each SLOT_EN read on a scope at or above 2.5 V throughout (the held high); then a MAIN tap and PI_KILL:
> every rail off, and at the next MAIN every SLOT_EN at 0 V before the panel runs".
<!-- /q -->

### A7. Stop conditions

- A supply at its limit in stage 1, or any input current over the stage's expected value by more than its stated tolerance.
- VBUS20 outside 19.08 to 20.96 V; VSYS under 12.054 V with no pack after EN_OOA 0; any rail outside Appendix A's tolerance or this
  page's band; a rail that is up with its enable off.
- A slot rail, PoE, the PA rail or an outlet rising before its enable is written; any SLOT_EN line above 0.266 V before the panel
  drives it.
- U42's limit acting (VSYS_DOCK collapsing) with nothing on pin 1; U44's or U45's limit acting at no load.
- **On a board without the VBUS20 cut: VIN_RAW over 24 V, ever.**
- A pack, or a stiff source, on CELL+ before TP-E11-30 has passed or Nexperia's acceptance is filed (R-160).
- A part heating with no load to explain it.

## Board B
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

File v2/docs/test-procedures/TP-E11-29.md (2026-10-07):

# TP-E11-29: the three battery FETs' installed thermal path and junction limit (Q39, Q40 and Q42)

<!-- tp
id: TP-E11-29
title: The three battery FETs' installed thermal path and junction limit (Q39, Q40 and Q42)
register: R-159
e11: E11-29
route5d: E11-29 (R-159)
-->

**Status: PROPOSED, for the supplier to review and agree before execution.** MESHSAT-1357, 3 October 2026; rewritten on 4 October
2026 on L4-E11's round 13 (its section 23), after the owner's supplier-delta review of that day (finding DELTA-02); its fixture and pass
rules rewritten on 5 October 2026 on L4-E11's round 14 (its section 24), after the independent recheck V2R, and its heavy leads, interlock,
galvanic boundary, SW_S's clamp, uncertainty and design target on round 15 (its section 25), after the final recheck V2RF; its heavy
leads restated as a requirement on the supplier's fixture on round 16 (its section 26), after the check V2RG. Prototype
design: nothing here has been built, bought, powered or measured. Common rules (the verdict rule, the record to keep, common safety):
`v2/docs/test-procedures/README.md`.

**NOT EXECUTABLE.** Two things must happen first: (1) the limits agreed: L4-E11's row E11-29 as section 8 quotes it, and the register's
row R-159 restated from it (L4-E9's), a restatement set 31 made word for word on the set 30 candidate and section 8 quotes since 6
October 2026, so this condition holds once the integration after set 30 (`fnd/int31regen`), which adopts this page's restated condition (set 30's promoted `dd1aed00` carries the re-quoted cells but its condition (1) still reads that the two quotes differ) is promoted and the checker's output is re-taken on it; (2)
a supplier's written agreement to the setup of section 5 (the fixture, its requirement on the heavy leads, and the coupon with its three
gates brought out apart). The checks so far, all AI reviews: the independent check V2R confirmed method (B) as an electrical method,
CONDITIONAL; the final recheck V2RF closed the fixture and the pass rules (V2R-B1, V2R-B2) AS CONDITIONAL and found round 14's
heavy-lead treatment unworkable (V2RF-B1); the check V2RG closed the interlock and V2RF's minors AS CONDITIONAL and found round 15's
guard NOT CLOSED (V2RG-B1), which ended the lead treatment's design loop. **With that, this procedure is ready to be PUT to a supplier
for agreement, the fixture requirement on the heavy leads (section 5, item 10) being the supplier's scope; V2RG-B1 stays OPEN as that
supplier qualification item** until the supplier's demonstration (step 0) shows the requirement met. The status line is in section 8.
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

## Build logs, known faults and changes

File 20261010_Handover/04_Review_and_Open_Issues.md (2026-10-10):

# Final review of Layers 1 to 3 and the open issues (handover of 10 October 2026)

**Scope of this review.** A bounded final read (about 30 minutes) by the coordinating agent session, from existing
evidence:
- Layer 1: purpose, users, scope and exclusions.
- Layer 2: scenarios, modes, interactions and the environment.
- Layer 3: identifiable requirements, acceptance criteria and traceability.
- Contradictions, missing files, broken links and later owner rulings.

It is an AI check, not a qualified engineering review. It re-uses the acceptance evidence named in `00_START_HERE.md`; it
does not repeat it. No requirement was changed and no source document was edited for this handover.

## 1. Findings on the baseline itself

- **Present and identifiable:**
  - Purpose, users, prototype scope and exclusions are stated (Layer 1 acceptance items 1.1 to 1.12, `LAYER-STATUS.md`).
  - The normal, degraded, startup, charging, shutdown, storage, service and fault scenarios, the envelope and the modes are stated (Layer 2 items 2.1 to 2.17).
  - Every requirement record has an identifier, a source link, an acceptance criterion where one is defined, an allocation, and a verification method and phase (Layer 3 items 3.1 to 3.18). `REQUIREMENTS-TRACE.md` carries the trace.
  - REQ-072 (runtime) is the registry's only design objective; every other record is mandatory.
- **Links:** every markdown link of the supplied core documents resolves inside this folder (checked by script at packaging). Citations written as repository paths in backticks are not links and resolve in the repository at the source commit.
- **Missing files:** none of the files the requirement pages link to is missing at the source commit.

## 2. Material issues

Kind: **INFO** = missing information or a record not yet updated; **FAIL** = an established design shortfall or failure
against a valid requirement; **PKG** = a packaging limitation of this handover.

| ID | Kind | Source | Affected | Practical consequence | Next engineering action |
|---|---|---|---|---|---|
| I-01 | INFO | `DEFINITION-CHANGE-RECORD-L3.md`; closure item L3-C63 | `PRODUCT-BRIEF.md`, `CONOPS.md` | The baselined texts still predate the owner's Layer 3 rulings D-32 to D-37; the change record governs where they differ (amendment A-2) | Write the change record's texts into both documents (re-stamp), keeping the accepted baselines as history |
| I-02 | INFO | `03_Requirements/APPROVED-AMENDMENTS.md` A-1 | D-06, D-01; `l3r2.yaml`, `REQUIREMENTS-L3-R2.md`, the definition texts | The second pack is approved (two identical, interchangeable complete 4S3P packs in the unchanged Peli 1450) but the registry and texts still read "D-06's one pack" | Add the approval to the registry as an amendment of D-06 with its exact scope; treat the one-pack restriction as superseded |
| I-03 | INFO | `REQUIREMENTS-L3-R2.md` section 2.6, rendered from `l3r2.yaml` (the `statuses` list) | the page's status table | It still reads the Layer 3 baseline "DRAFTED ... Not yet validated and accepted", although `baseline_acceptance` records acceptance at `3b4b92cf` (and `LAYER-STATUS.md` agrees). Editing it here would break the registry's content-bound acceptance | Read `baseline_acceptance` as governing; correct the status entry at the next registry revision and re-render |
| I-04 | FAIL (objective) | record l4rt (fnd/l4rt `3964c68a`), its two-pack coverage (fnd/l4rt72 `667c297e`, checked W360/W362); MODEL figures | REQ-072, 48 to 72 h at PS-IDLE-SPEC (42.8 W) | One pack runs about 2.5 h on battery; two packs about 5.04 h at +20 C and 2.08 h at -10 C; a September night is short by about 255 Wh; all 42 full-service rows FAIL (December 46 of 46). Only a reduced night mode (not approved; as drawn it hosts neither Iridium nor the SOS path) reaches zero, at +20 C only. The bus-voltage basis is the model's most favourable (feasibility finding F-01) | Keep REQ-072 as written; the runtime against service is the owner's scope question (section 3) |
| I-05 | FAIL | `REQUIREMENTS-L3-R2.md` 2.6 (DR-02, DR-03); Layer 4 records | power path, outlet contracts | Board A's power path as drawn fails (DR-02) and the outlet trips below its contracts (DR-03); Layer 4's desk gate is not passed and power closure is blocked | Re-architect or correct the power path in Layer 4 against the requirements |
| I-06 | FAIL (coverage) + INFO | record l4e12 section 21 (fnd/l4cfl `1eaf9d55`, checked W363 then W366) | REQ-042 battery-bay VOC sensing (CHO-001, SC-41) | The SGP41 covers VOC only to +50 C against bay air up to about 70 C. A Layer 4 working selection adds the Honeywell BES Series (-40 to +85 C, 0 to 90 %RH), CONDITIONAL: no printed trip concentration or maximum current, its bay fit, its CAN interface and the closed-bay test are open, and its maker states it is not a safety or emergency stop device | Verify the selection's conditions; answer the safety-device question (section 3) |
| I-07 | INFO | record l4e12 (closed-lid thermal arrangement), U-02, T-H1 | thermal requirements | The closed-lid arrangement is conditional on a physical thermal test (T-H1) that has not run | Run or commission T-H1 before thermal closure |
| I-08 | INFO | U-01 (bench E-01); record l4pk2; appendix 32.62 vs the pocket-fit check | cells, pack fit | Cell suitability is unqualified; the second pack's fit is unproven; the buildable store is recorded as 268.9 Wh in one source and 215.8 Wh in another | Qualify the cell; resolve the volume conflict from the case model; prove the two-pack fit |
| I-09 | FAIL (drafted fixes) | records l4checkb, l4emc (checked W373/W376), l4seat | board B EMCON lines; layout entry | Three EMCON circuit defects (U544 in fault F6, U543's pull-up, RB_IEN during U543's reset delay) have drafted corrections, unapplied. A further window (RB_IEN while +5V_DEV is under 2.6 V) is open. Board B's seating is incomplete (the last placed board had 6 hard violations and 178 decoupling-distance failures) | Apply or redesign in the board B round; do not start layout before it places clean |
| I-10 | PKG | repository state | Layer 4 working material | The unintegrated Layer 4 branches exist only in the programme's runner repository (not published) | Request the bundle named in `05_Engineer_Takeover.md` if that material is wanted |
| I-11 | PKG | all acceptance records | Layers 1 to 3 | Every acceptance rests on AI reviews and AI checks; none is a qualified engineering review | Hold the engineer's own review of the baseline as part of the takeover |

## 3. Product-scope questions (for the owner; they do not block the takeover)

1. **REQ-072, runtime against service.** No studied configuration meets 48 h at full service, including the approved two packs. The routes on record each reopen an owner ruling:
   - accept the shortfall (excluded by D-20 as recorded);
   - a reduced night mode, which turns services off;
   - a larger store, which is limited by the unchanged case.

   The record's plain-language restatement is in fnd/l4rt72 `L4RT.md` section 9.4.
2. **REQ-042, the gas shutdown's safety basis.** Whether the battery-bay gas shutdown needs a rated safety device. Both sensor makers disclaim safety use; the pack's own hardware protection does not depend on either sensor.

Routine technical choices (copper, stackup, components, routing, methods, test setups) are the receiving engineer's and are not listed here.

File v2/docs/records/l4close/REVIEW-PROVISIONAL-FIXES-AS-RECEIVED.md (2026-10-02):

# MeshSat Layer 4: review of the provisional power fixes

**Review date:** 2 October 2026  
**Reviewed:** rejected candidate `8fbb68b6`, correction packet at `516d43fe`, and separate B6 addendum at `11339ec7`.  
**Verdict:** useful corrections, but **B2 and B6 are not demonstrated closed**. B1's supply reroute also needs a branch-fault protection decision. This is an engineering review of supplied drafts, not fabrication approval.

The immediate work is now specific: qualify the battery switch, give the solar guard a defensible component and interconnect envelope, and protect the new auxiliary feed. The charging-loss correction is sound. The runtime correction properly separates energy-only endurance from service reduced by temperature. Preserve those results.

## 1. What I actually reviewed

| Input | Bytes | SHA-256 | Manifest result |
|---|---:|---|---|
| `MESHSAT-L4-POWER-PACKET-PREVIEW-8fbb68b6.zip` | 6,388,336 | `b2cf128e913e1f2eb3a4e03d6a041678c87d50ffa41035814af75c304b490786` | 340 entries, all match |
| `MESHSAT-L4-PROVISIONAL-FIX-REVIEW-8fbb68b6-to-516d43fe.zip` | 1,509,068 | `c1ac471462259596d76ec192a8b8ad8ea70ddec8f982546ccad8f8aa64fe8bb9` | 36 entries, all match |
| `MESHSAT-L4-PROVISIONAL-FIX-REVIEW-ADDENDUM-B6-11339ec7.zip` | 290,980 | `c2a8c77d89dbc4114d6599f73c34b80be776d459e4939d61a8de20dc0ae22f45` | 8 entries, all match |

I read Astra's seven-blocker report, the changed calculations, draft circuit edits, affected tests and consolidated claims. I independently recomputed selected electrical and thermal results and exercised the B6 numerical function in a separate sensitivity harness.

I applied the audited constant edit tables **in memory**, against the supplied generator text: board A's 16 edits, board E's 17 edits and the interface YAML's five edits apply and parse. The target `check_contracts.py` is absent, so its alias edit was not exercised. All **15 changed Python files** parse successfully. These checks establish neither circuit correctness nor a passing integrated suite.

The inspection overlay is not a real Git revision. I did not execute the complete project test suite, bypass source-hash gates, run KiCad, modify the design, or test hardware. Manufacturer PDFs are largely omitted. I separately retrieved the official Nexperia FET and TI charger documentation. The Saft portal's direct PDF open failed; the B5 assessment below therefore concerns the corrected qualification claim, not an independently completed cell qualification.

**Not reviewed:** subsequently reported integration `c0916a6c`, the final merged B6 candidate, and its targeted Astra recheck. A coordinator's status report is not evidence that those revisions pass this review.

## 2. Disposition of Astra's seven blockers

“Corrected” below means the identified error is corrected within this review's stated scope. It does not mean the proposed hardware has been implemented or qualified.

| Blocker | Disposition | Basis and remaining obligation |
|---|---|---|
| **B1 — E's auxiliary feed and startup claim** | **Topology corrected; qualification open** | U12, its input capacitor and the fans move to VSYS through coordinated A/E dock edits. The unsupported startup-time guarantee is withdrawn. Successful source-only startup and held-pack drain remain conditional. New branch protection gap: L4-F03 below. |
| **B2 — battery FET** | **Not closed** | Replacement is a candidate, but the proposed thermal and body-diode qualifications rely on assumptions not covered by the stated closing tests. See L4-F02. |
| **B3 — thermal modes and limits** | **Substantially corrected; classification needs correction** | Local limits and the SGP41 sensing limit are distinguished. However, the consolidation still turns model-dependent ceilings and missing e-paper storage evidence into physical impossibility and owner conflicts. See L4-F04. |
| **B4 — charging heat** | **Arithmetic correction accepted** | Independently obtained 50.04366 W, or 52.13366 W including the stated ballasts. This validates the correction under the stated inputs; it does not qualify those inputs or the enclosure. |
| **B5 — Saft current-versus-temperature claim** | **Overclaim corrected** | Current at temperature, dwell/recovery and fit now remain open explicitly. Approval to adopt the cell and physical qualification remain outstanding. |
| **B6 — guard already on during a fault** | **Not closed** | A real transient model now exists, but cable inductance alone is insufficient to qualify it. Capacitor assumptions and model uncertainty matter at the very small margin. See L4-F01. |
| **B7 — battery runtime versus thermal response** | **Original reasoning error corrected** | The 2.52 h value is labelled energy-only; the model now includes load shedding. I reproduced the constant-conductance counterexample. The nonlinear enclosure and actual hardware temperatures remain unqualified. |

## 3. Findings requiring action

### L4-F01 — P1: B6's stated cable condition does not establish a robust transient bound

**Evidence:** B6 version of `v2/docs/records/l4e7/l4e7_stage_settings.py`, lines 215–324, 1898, 2383, 2505–2519, 2527–2597 and 2671–2673; its output, lines 869–965; `test_l4e7.py`, lines 827–866.

The supplied result is **0.2991 V against U5's 0.3000 V absolute limit**, conditional on at least **2.47 µH** in the panel lead. That is approximately **0.9 mV, or 0.3%, headroom**.

The code uses one bias factor `k` for three capacitor banks: the ceramics on PV_P, those on TRK_VS, and C13/C14 on TRK_VIN. The banks' initial tolerances are treated separately, but their uncertain DC-bias behaviour is tied together. No manufacturer's part/curve establishes that correlation. Other assumptions include a 0.25 bias floor for the 100 V port capacitors and 10 mΩ ceramic ESR.

I reconstructed the worst reported operating case from printed values and formulas: 36 V source step, 7.46 V initial state, no initial load, 2.47 µH lead, aged cold bulk. This is a **rounded-input reconstruction, not an exact replay of the complete generator**.

| Numerical check | U5 positive sense differential |
|---|---:|
| Supplied function, reconstructed inputs, 20 ns timestep | 0.299128 V |
| Same inputs, 1 ns timestep | 0.299598 V |
| 20 ns, TRK_VS bias factor 0.99, downstream factor 1.00; other factors unchanged | **0.300218 V** |
| 20 ns, TRK_VS bias factor 0.95, downstream factor 1.00 | **0.304662 V** |

The finer timestep alone does **not** prove failure; it consumes about half the original margin. The independent-factor checks are sensitivities, not a claim that a particular purchased capacitor has these characteristics. Their significance is that the current evidence does not exclude them. **Meeting the lead-inductance condition therefore does not, by itself, establish the rating claim.**

The current numerical test usefully checks a simplified RLC response, but allows 1% peak error in that test. It does not establish error below this design's approximately 0.3% sense-voltage margin in the switched, loaded network.

**Required correction:** select actual capacitors and bound effective capacitance, ESR and relevant parasitics at their respective voltages and temperatures. Separate bank parameters unless correlation is supported. Include numerical error in the margin. Specify the complete permissible lead/source/fault-location envelope; a theoretical spacing calculation is not a measured harness specification. If protection requires minimum inductance, make it a controlled, toleranced part of the design or qualify the complete constrained harness. Do not assume every fault traverses five metres of lead.

**Closure:** the selected network must meet the ratings with explicit margin over its bounded uncertainties and the declared fault envelope. Reproduce the critical cases independently and confirm the subsequent bench waveforms at the IC pins. If this topology cannot provide margin, change the protection network rather than repeatedly searching for the smallest passing cable inductance. Preserve the valid corrections to CS115's interpretation.

### L4-F02 — P1: B2's replacement FET qualification still overstates what is established

**Evidence:** `v2/docs/records/l4e11/l4e11_power.py`, lines 2213–2226, 2305–2308, 2321–2339, 2350–2380 and 2468–2514; output rows E11-29/E11-30; `test_l4e11.py`, lines 762–786.

The two BUK6Y10-30P devices may be a workable selection. The supplied proof does not yet demonstrate that:

- `fet_bound()` assumes convex interpolation and a temperature-independent upper bound on the gate-voltage ratio. It produces **21.136 mΩ at 8.5 V and 150 °C**, explicitly through inference. That is not a printed maximum at the operating point.
- The transient thermal shape comes from **the previous AOS device**, scaled for the new devices. A case-rise measurement at 10 A cannot establish that borrowed transient shape for all the listed fault pulses. Adjacent devices' thermal coupling also needs an explicit treatment.
- The code treats **4.72 nF of typical capacitance** as meeting the 5 nF selection criterion without establishing the required margin over operating conditions and variation.
- The docking check converts a **320 A, ≤10 µs pulse rating** into **1.024 A²s**, then accepts an exponential pulse with a **33.8 µs time constant** because its calculated I²t is smaller. The source does not provide that I²t rating. Matching diode paths alone does not validate the conversion or the assumed hot derating.

The official [Nexperia BUK6Y10-30P sheet](https://assets.nexperia.com/documents/data-sheet/BUK6Y10-30P.pdf), pp. 2–6, gives resistance maxima at specified test points, a typical capacitance, and the stated short pulse condition. [TI's BQ25730 sheet](https://www.ti.com/lit/ds/symlink/bq25730.pdf), p. 92, recommends P-channel BATFET input capacitance below 5 nF. These support the distinction between a candidate selection and completed qualification. Nexperia's [thermal/current application note](https://assets.nexperia.com/documents/application-note/AN90016.pdf) also distinguishes steady thermal resistance from transient impedance and relates body-diode loss to voltage times current; it is not authorization for this pulse extrapolation.

**Required correction:** use a device-specific electrothermal/qualification basis with justified uncertainty and margin. Check the actual 18 A/60 s service and relevant fault histories from the hot initial state. Qualify the complete diode-inrush waveform and sharing, or constrain that waveform through precharge/current limiting. If a different switch gives a simpler supported design, choose it. Do not lower the required service to make the part pass.

**Closure:** updated analysis and tests address the assumptions actually used. E11-29's steady case-rise check and E11-30's sharing check alone are insufficient. This finding establishes a qualification gap, **not a demonstrated physical failure of the replacement FETs**.

### L4-F03 — P1: the new VSYS_E contact needs branch-fault protection

**Evidence:** `apply_gen_sch_a_charger.py`, lines 79–89; `apply_gen_sch_e_aux.py`, lines 35–66; `apply_pcb_interfaces_dock.py`, lines 31–50, all under `v2/docs/records/l4e11/`.

Moving E's auxiliary load to VSYS fixes the original supply-path error. The draft connects the high-current VSYS rail directly to **one dock contact rated in the record at 3.5 A**. The 1 A load declaration is bookkeeping, not a current limiter. No branch fuse or current-limiting element is introduced in these edits.

The common power path is designed for 10 A continuous and 18 A pulses, with much higher upstream protection thresholds. That does not establish protection of this smaller branch. A concrete analysis case is an overload drawing 5 A from 14.4 V—equivalent to 2.88 Ω—on VSYS_E: above the contact's stated rating but below the source path's declared continuous capability. This is an electrical counterexample to relying on the 1 A declaration, not a claim that the built connector has already failed.

**Required correction:** bound this branch's overload, short-circuit, inrush and recovery currents, including source-only and battery operation. Add coordinated branch protection or demonstrate another physical limiting mechanism that protects the contact, wiring and copper over temperature and the required pulse durations. Check the new feed's voltage drop against E's startup and fan requirements.

The old cross-board supply topology need not be reopened. Complete this local protection design as part of the coordinated A/E/interface patch.

**Related claim to correct:** `L4-POWER-ARCHITECTURE.md` around line 821 says the held-pack drains are bounded at 0.1408 mA. The underlying L4-E11 section 15a explicitly leaves hot clamp leakage and body-diode current unbounded. Describe 0.1408 mA as the quantified subset, and preserve the separate ≤1 mA bench acceptance.

### L4-F04 — P2: thermal screening is being promoted into proof of impossibility

**Evidence:** `v2/docs/records/l4e12/l4e12_thermal.py`, `govern()` around lines 539–565, `per_mode()` lines 1831–1882, and `caps()` lines 2027–2075; output section 12e; correction packet's `BLOCKER-DISPOSITION.md`, B3.

The corrected mode table is useful. The subsequent claim that four rows “exceed any measurable capacity” is too strong:

- The e-paper has no held unpowered-storage limit. Using its operating limit as a conservative screening assumption does not prove that an unpowered device cannot survive a higher temperature.
- The capacity comparison uses chosen convection/radiation coefficients and particular heat paths. An optimistic model endpoint is not automatically a demonstrated upper bound on every compliant physical implementation.
- The addendum itself identifies a local e-paper temperature measurement and a closed-lid conduction route that could change the outcome. That contradicts an unconditional “no measurement can pass” summary.

**Required correction:** distinguish **modelled failure of the analysed arrangement**, **missing storage qualification**, and **a demonstrated conflict with mandatory requirements**. Keep local part temperatures separate from mixed-air screens. Only the last category justifies asking the owner to weaken a requirement; the other two remain bounded engineering or evidence tasks.

This does not establish that the sealed case will work. T-H1 and the applicable local temperature/storage evidence remain necessary. It prevents an unsupported impossibility claim from forcing another owner-decision loop.

## 4. Results worth preserving

**B4 — charging heat.** With the supplied load 42.82355 W, 46.5 W into the pack, combined efficiency 0.95 × 0.98 and 0.6 W cell loss:

`P_input = (42.82355 + 46.5) / (0.95 × 0.98) = 95.943663 W`

`P_stored = 46.5 − 0.6 = 45.9 W`

`Q_case = 95.943663 − 45.9 = 50.043663 W`

Adding the stated 2.09 W ballast allowance gives **52.133663 W**. This agrees with the correction. The previously omitted load-supply loss is **3.173818 W**. Do not reopen this arithmetic unless the topology, loads, efficiency basis or thermal boundary changes.

**B7 — thermal response.** At 43.413 W case heat, 0.6711 W/K conductance, 8 kJ/K thermal mass and a +20 °C start, the closed-form model reaches +50 °C after **2.06349 h**. Without shedding it reaches **54.467 °C at 2.52 h**. A runtime shorter than the time constant was never sufficient to exempt thermal limits. The revised text fixes that reasoning. Its reported 2.52–2.95 h after shedding must remain distinguishable from uninterrupted operation at the original profile.

**B5 — cell selection.** The corrected report explicitly says the proposed Saft cell's temperature window does not prove simultaneous current/temperature capability, dwell recovery or fit. Keep that qualification. Its energy comparison borrows Samsung discharge-curve behaviour, so treat the Saft runtime numbers as sensitivities until cell-specific evidence replaces them. This neither authorizes a cell purchase nor changes the owner's approved pack arrangement.

**B1 — coordinated edits.** The A/E/interface changes address the original pack-side-feed mistake. Preserve that topology while resolving L4-F03, startup qualification, fan voltage rating and held-pack current.

## 5. A bounded path forward

Keep the accepted Layer 3 requirements baseline. The runtime objective remains a reported design shortfall; it is not a reason to restart requirements work.

Within the existing two-worker limit:

1. One electrical author closes **B2 and the new auxiliary-feed protection**, using the actual combined A/E draft.
2. One electrical author closes **B6's component, lead and transient envelope**, starting from the supplied sensitivity witnesses. Decide the intended margin before selecting values.
3. Correct the thermal classifications in the existing consolidation. Do not commission another broad thermal review merely to restate the same uncertainty.
4. Give Astra the resulting **exact integrated commit**, the four findings here, and the decision-critical calculations. Its check should challenge the selected assumptions and physical margins, not only reproduce script output. Preserve independently confirmed corrections.
5. Maintain separate outcomes: **reviewed architecture**, **implemented circuit**, and **prototype qualification**. A condition with a named owner and test is useful handover material; it is not evidence the condition has passed. Reviewer run limits also do not turn an unresolved finding into acceptance.

If a supported solution remains unavailable, deliver the connected design and these narrowly defined open items to the electronics engineer now. Do not delay that handover to polish every generated page. A useful engineer packet consists of the proposed circuit changes, operating/fault envelope, calculations, unresolved assumptions and exact acceptance tests.

**What this review does not justify:** “power solved,” “Layer 4 100% complete,” or a new completion ETA. It does justify retaining the corrected B4 arithmetic, B7 reasoning and B5 qualification language while directing the remaining work at specific electrical decisions.

## 6. Reproduction companion

`meshsat-layer4-review-checks-2026-10-02.zip` contains the extracted pure `guard_event` function, sensitivity probes, arithmetic/draft-check harness, machine-readable results and provenance. The B6 probes run independently of the repository; the draft checks require the supplied packet overlay. No acceptance guard is removed.

The numerical witness uses printed, sometimes rounded, input values. Its baseline agrees with the reported sense differential to the printed four decimal places. It demonstrates fragility and missing parameter coverage, not a completed SPICE/bench validation or an exact replay of the missing integrated candidate.

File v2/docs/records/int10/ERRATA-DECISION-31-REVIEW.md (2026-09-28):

# Erratum: the review of decision 31, the wall port eFuse's limit

MESHSAT-1357, integration set 9, stream s99reg, 29 September 2026. AI engineering work; prototype design, nothing
built, ordered or measured.

**Where:** `v2/docs/reviews/DECISION-31-PROTECTION-TOPOLOGY.md` line 244, the VBUS_WALL paragraph of board A's wall USB
host port: "VBUS_WALL is 5.0 V behind the eFuse U32 (limit 0.89 A)".

**Correction:** U32's limit is **0.9142 A nominal**. TPS2596 equation 7 (TI SLVSET8A, May 2019, revised August 2019,
printed p.28) is RILM = 903 / (ILIM - 0.0112); the page's worked example, 903 / (1 - 0.0112) = 913.2 ohm, fixes the
sign. With R186 at 1.00 kOhm, ILIM = 903 / 1000 + 0.0112 = 0.9142 A. The 0.89 A came from the generator's comment,
which carried the sign as + (stream s99a corrected the generator, `v2/docs/records/s99a/README.md` section 2; the
independent check of s99a reproduced it). No maximum at 1 kOhm is published: the 909 ohm row of SLVSET8A p.6 scaled to
1 kOhm gives about 0.956 A, an estimate.

**What the correction changes in the review:** nothing it concludes. The paragraph reads the ESD array's clamping
voltage against U32's output rating and C156's hold-up in a discharge; the limit is quoted as context and enters no
figure of the paragraph (0.055 V at 8 kV and 0.10 V at 15 kV are C156's, independent of the limit).

**Why the review is not edited:** its sha256 (`0948170232...`) is pinned three times in `v2/ecad/tools/pcb_board_holds.yaml`,
as the review requirement of the holds of boards A, D and E, and the reviewed port set cites the review. Editing it
turns each hold's review requirement to "re-review it", and the pinning script
(`v2/docs/records/d8dec31/apply_holds_review_pin.py`) cannot re-pin: it refuses unless the netlists in the tree are the
ones the review read (board A's has moved since, and moves again with decision 55's regeneration). The review stays as
filed; `v2/docs/records/int10/apply_pages_s99.py` asserts it is byte-identical to its pins and that this erratum is
present. Any later review of board A should quote 0.9142 A; none is owed by the regeneration itself, since the decision 31 hold's review pin moved to the new netlist on a parsed proof and reads met (set 9's AI check, minor item M4).

**Other places the wrong-sign figure stays, as history (not edited):** `v2/docs/records/r4a/r4-decisions.md` line 196
("ILM 1.00 k = 0.89 A") and `v2/docs/records/r4b/r4-interfaces.md` line 11 (records of round 4 streams), and the frozen
handover snapshot `v2/release/handover/H1/` (its copies of `gen_sch_a.py`, `pcb_interfaces.yaml`, `ASSEMBLY.md` and the
two records). Each reads 0.9142 A nominal by this erratum. The live pages are corrected by
`v2/docs/records/int10/apply_pages_s99.py` (HW-FW-CONTRACT.md FW-A07, ASSEMBLY.md section 4) and
`apply_if_ab_power_s99.py` (pcb_interfaces.yaml IF-AB-WALL).

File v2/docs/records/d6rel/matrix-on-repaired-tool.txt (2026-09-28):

THE FOUR-CASE MATRIX ON THE REPAIRED TOOL (worker d6rel, MESHSAT-1357, taken 28 September 2026 17:55 CEST, after the fixes of the fresh check: a class whose maker publishes no figure holds its board, every open item holds a reading, jack, RJ45 and plug in the word net)
The tool is v2/ecad/tools/reliability.py of this branch; case 4's list is v2/ecad/tools/pcb_reliability.yaml beside it, whole, asked for board A. Command, from the worktree root:
  python3 v2/docs/records/d6rel/matrix.py v2/ecad/tools v2/ecad/tools/reliability.py
Exit code of the matrix script: 0 (the four cases read PASS, FAIL, FAIL, INCONCLUSIVE, as the review asks). The fixture sheets of cases 1 to 3 are pinned to the fixture netlist's sha by matrix.py; their one class cites its figure, so case 1 may read PASS.
Nothing was built or measured: these are readings of fixture netlists.

tool under test : <worktree>/v2/ecad/tools/reliability.py  sha256/16 c50f2b8b35d1d57b
tools directory : <worktree>/v2/ecad/tools
case 4's list   : <worktree>/v2/ecad/tools/pcb_reliability.yaml  sha256/16 40f2a98323b1f9ce
fixtures in     : a temporary directory outside the tree (mkdtemp prefix d6rel-matrix-)

== case 1-one-declared-jst: one declared JST connector
   wanted PASS (exit 0); the tool says PASS (exit 0): as wanted
   counts {"boards": 1, "candidates": 1, "citations_unjudged": 0, "classed": 1, "classes": 1, "classes_undecided": 0, "covered": 1, "excluded": 0, "exclusions": 0, "fail": 0, "figures_cited": 1, "figures_none_published": 0, "figures_not_mated": 0, "figures_owed": 0, "inconclusive": 0, "measures_owed": 0, "per_board": {"a": {"artefact": {"kind": "netlist", "sha256_16": "ed25c2105c339c38"}, "bound": true, "candidates": 1, "citations_unjudged": 0, "classed": 1, "classes_undecided": 0, "excluded": 0, "held_by": [], "refused": 0, "result": "PASS"}}, "refused": 0}  denominator 1  missing_input None
   inputs recorded: {"board": "a", "list": {"path": "<fixtures>/1-one-declared-jst/list.yaml", "sha256": "d7e72f12592c2343ff26dc04e17b6c6fe8a9245a16ebd84a92914d6a3de0b3d9", "sha256_16": "d7e72f12592c2343"}, "netlist": {"content16": "8649156fa63ebb2d", "parts": 1, "path": "<fixtures>/1-one-declared-jst/ecad/pcb-a-power/out/pcb-a-power.net", "sha256": "ed25c2105c339c38025ded5885383f2ff5ab3f65eb9107b3ffeb133e27418620", "sha256_16": "ed25c2105c339c38"}}
   | reliability: the list <fixtures>/1-one-declared-jst/list.yaml sha256 d7e72f12592c2343ff26dc04e17b6c6fe8a9245a16ebd84a92914d6a3de0b3d9
   | reliability: A   PASS         netlist <fixtures>/1-one-declared-jst/ecad/pcb-a-power/out/pcb-a-power.net sha256 ed25c2105c339c38025ded5885383f2ff5ab3f65eb9107b3ffeb133e27418620, 1 part(s)
   |              1 candidate(s): 1 classed in 1 class(es), 0 excluded by 0 exclusion(s), 0 refused; figures: 1 cited, 0 none published, 0 not mated, 0 owed; measures owed: 0
   | verdict: reliability            PASS         of 1 {"boards": 1, "candidates": 1, "citations_unjudged": 0, "classed": 1, "classes": 1, "classes_undecided": 0, "covered": 1, "excluded": 0, "exclusions": 0, "fail": 0, "figures_cited": 1, "figures_none_published": 0, "figures_not_mated": 0, "figures_owed": 0, "inconclusive": 0, "measures_owed": 0, "per_board": {"a": {"artefact": {"kind": "netlist", "sha256_16": "ed25c2105c339c38"}, "bound": true, "candidates": 1, "citations_unjudged": 0, "classed": 1, "classes_undecided": 0, "excluded": 0, "held_by": [], "refused": 0, "result": "PASS"}}, "refused": 0} | every candidate part of the inventory falls in one declared class, with its cycle figure from the maker's document or the reason it has none, its load and the measure taken, or under one declared exclusion with its reason. A desk reading of a netlist and a list: it tests nothing and replaces no physical verification; REL-001 is verified at the prototype and no board has been built

== case 2-plus-undeclared-idc: plus an undeclared IDC header
   wanted FAIL (exit 1); the tool says FAIL (exit 1): as wanted
   counts {"boards": 1, "candidates": 2, "citations_unjudged": 0, "classed": 1, "classes": 1, "classes_undecided": 0, "covered": 1, "excluded": 0, "exclusions": 0, "fail": 1, "figures_cited": 1, "figures_none_published": 0, "figures_not_mated": 0, "figures_owed": 0, "inconclusive": 0, "measures_owed": 0, "per_board": {"a": {"artefact": {"kind": "netlist", "sha256_16": "9e47827f307ef37d"}, "bound": true, "candidates": 2, "citations_unjudged": 0, "classed": 1, "classes_undecided": 0, "excluded": 0, "held_by": [], "refused": 1, "result": "FAIL"}}, "refused": 1}  denominator 2  missing_input None
   inputs recorded: {"board": "a", "list": {"path": "<fixtures>/2-plus-undeclared-idc/list.yaml", "sha256": "3c683a36c35b485b6e2d50c0228198a405f1a53a9018a77a37b525715d1cedb0", "sha256_16": "3c683a36c35b485b"}, "netlist": {"content16": "4526a971764f5144", "parts": 2, "path": "<fixtures>/2-plus-undeclared-idc/ecad/pcb-a-power/out/pcb-a-power.net", "sha256": "9e47827f307ef37d0300847ba0ae3debd658bc3a1300bb12ad5f0b8844d668ff", "sha256_16": "9e47827f307ef37d"}}
   | reliability: the list <fixtures>/2-plus-undeclared-idc/list.yaml sha256 3c683a36c35b485b6e2d50c0228198a405f1a53a9018a77a37b525715d1cedb0
   | reliability: A   FAIL         netlist <fixtures>/2-plus-undeclared-idc/ecad/pcb-a-power/out/pcb-a-power.net sha256 9e47827f307ef37d0300847ba0ae3debd658bc3a1300bb12ad5f0b8844d668ff, 2 part(s)
   |              2 candidate(s): 1 classed in 1 class(es), 0 excluded by 0 exclusion(s), 1 refused; figures: 1 cited, 0 none published, 0 not mated, 0 owed; measures owed: 0
   |   FAIL A: J_RIB1 (fixture ribbon (IDC 2x5)) carries load or sees cycling and is in no declared class and under no declared exclusion: reference class J (a connector)
   | verdict: reliability            FAIL         of 2 {"boards": 1, "candidates": 2, "citations_unjudged": 0, "classed": 1, "classes": 1, "classes_undecided": 0, "covered": 1, "excluded": 0, "exclusions": 0, "fail": 1, "figures_cited": 1, "figures_none_published": 0, "figures_not_mated": 0, "figures_owed": 0, "inconclusive": 0, "measures_owed": 0, "per_board": {"a": {"artefact": {"kind": "netlist", "sha256_16": "9e47827f307ef37d"}, "bound": true, "candidates": 2, "citations_unjudged": 0, "classed": 1, "classes_undecided": 0, "excluded": 0, "held_by": [], "refused": 1, "result": "FAIL"}}, "refused": 1} | every candidate part of the inventory falls in one declared class, with its cycle figure from the maker's document or the reason it has none, its load and the measure taken, or under one declared exclusion with its reason. A desk reading of a netlist and a list: it tests nothing and replaces no physical verification; REL-001 is verified at the prototype and no board has been built

== case 3-plus-undeclared-rj45: plus an undeclared "RJ45 MagJack"
   wanted FAIL (exit 1); the tool says FAIL (exit 1): as wanted
   counts {"boards": 1, "candidates": 2, "citations_unjudged": 0, "classed": 1, "classes": 1, "classes_undecided": 0, "covered": 1, "excluded": 0, "exclusions": 0, "fail": 1, "figures_cited": 1, "figures_none_published": 0, "figures_not_mated": 0, "figures_owed": 0, "inconclusive": 0, "measures_owed": 0, "per_board": {"a": {"artefact": {"kind": "netlist", "sha256_16": "575299cd4ce2143e"}, "bound": true, "candidates": 2, "citations_unjudged": 0, "classed": 1, "classes_undecided": 0, "excluded": 0, "held_by": [], "refused": 1, "result": "FAIL"}}, "refused": 1}  denominator 2  missing_input None
   inputs recorded: {"board": "a", "list": {"path": "<fixtures>/3-plus-undeclared-rj45/list.yaml", "sha256": "646353cb9f3a5f9015ae1bc24134da42b675c20ddac818d62b5b9163aef51b30", "sha256_16": "646353cb9f3a5f90"}, "netlist": {"content16": "5f0494a7619fc4c8", "parts": 2, "path": "<fixtures>/3-plus-undeclared-rj45/ecad/pcb-a-power/out/pcb-a-power.net", "sha256": "575299cd4ce2143e1e8d23801211aeb9fc864f85c959b36fb3f32373ca90dea7", "sha256_16": "575299cd4ce2143e"}}
   | reliability: the list <fixtures>/3-plus-undeclared-rj45/list.yaml sha256 646353cb9f3a5f9015ae1bc24134da42b675c20ddac818d62b5b9163aef51b30
   | reliability: A   FAIL         netlist <fixtures>/3-plus-undeclared-rj45/ecad/pcb-a-power/out/pcb-a-power.net sha256 575299cd4ce2143e1e8d23801211aeb9fc864f85c959b36fb3f32373ca90dea7, 2 part(s)
   |              2 candidate(s): 1 classed in 1 class(es), 0 excluded by 0 exclusion(s), 1 refused; figures: 1 cited, 0 none published, 0 not mated, 0 owed; measures owed: 0
   |   FAIL A: J_ETH (RJ45 MagJack) carries load or sees cycling and is in no declared class and under no declared exclusion: reference class J (a connector)
   | verdict: reliability            FAIL         of 2 {"boards": 1, "candidates": 2, "citations_unjudged": 0, "classed": 1, "classes": 1, "classes_undecided": 0, "covered": 1, "excluded": 0, "exclusions": 0, "fail": 1, "figures_cited": 1, "figures_none_published": 0, "figures_not_mated": 0, "figures_owed": 0, "inconclusive": 0, "measures_owed": 0, "per_board": {"a": {"artefact": {"kind": "netlist", "sha256_16": "575299cd4ce2143e"}, "bound": true, "candidates": 2, "citations_unjudged": 0, "classed": 1, "classes_undecided": 0, "excluded": 0, "held_by": [], "refused": 1, "result": "FAIL"}}, "refused": 1} | every candidate part of the inventory falls in one declared class, with its cycle figure from the maker's document or the reason it has none, its load and the measure taken, or under one declared exclusion with its reason. A desk reading of a netlist and a list: it tests nothing and replaces no physical verification; REL-001 is verified at the prototype and no board has been built

== case 4-board-a-no-netlist: board A's declaration and no netlist
   wanted INCONCLUSIVE (exit 3); the tool says INCONCLUSIVE (exit 3): as wanted
   counts {"boards": 1, "candidates": 0, "citations_unjudged": 0, "classed": 0, "classes": 11, "classes_undecided": 4, "covered": 0, "excluded": 0, "exclusions": 1, "fail": 0, "figures_cited": 5, "figures_none_published": 4, "figures_not_mated": 0, "figures_owed": 2, "inconclusive": 10, "measures_owed": 0, "per_board": {"a": {"artefact": null, "bound": false, "candidates": 0, "citations_unjudged": 0, "classed": 0, "classes_undecided": 4, "excluded": 0, "held_by": ["REL-O-01", "REL-O-02", "REL-O-07", "REL-O-08", "REL-O-12", "REL-O-13"], "refused": 0, "result": "INCONCLUSIVE"}}, "refused": 0}  denominator 0  missing_input 'board A has no netlist of its declared phase in this tree (/tmp/d6rel-matrix-glndel24/4-board-a-no-netlist/ecad/pcb-a-power/out/pcb-a-power.net)'
   inputs recorded: {"board": "a", "list": {"path": "<fixtures>/4-board-a-no-netlist/list.yaml", "sha256": "40f2a98323b1f9ceeea024fac42b46521d565f0547ee6824ff29dcd5ddaabd96", "sha256_16": "40f2a98323b1f9ce"}}
   | reliability: the list <fixtures>/4-board-a-no-netlist/list.yaml sha256 40f2a98323b1f9ceeea024fac42b46521d565f0547ee6824ff29dcd5ddaabd96
   | reliability: A   INCONCLUSIVE no artefact read
   |   note board A has no netlist of its declared phase in this tree (<fixtures>/4-board-a-no-netlist/ecad/pcb-a-power/out/pcb-a-power.net), so the list could not be compared with the board
   |   INCONCLUSIVE board A has no netlist of its declared phase in this tree (<fixtures>/4-board-a-no-netlist/ecad/pcb-a-power/out/pcb-a-power.net)
   |   INCONCLUSIVE A: class the pre-charge pin owes its cycle figure (open item REL-O-01: board A's pre-charge pin J_PRE1, the longer Mill-Max pin that mates first, has no order code: its value in the netlist names no part ('pre-charge pin, longer, mates first (32.24 AX)') and no document of a longer pin is held, so no maker's figure can be cited for it)
   |   INCONCLUSIVE A: class the USB-C outlet's pigtail header owes its cycle figure (open item REL-O-02: the 2.54 mm pin header lands carry no named part: their values in the netlists name the lead, the module or the bench use and no header, and whether a header is fitted or the lead is soldered into the holes is a build choice not made. ASSEMBLY.md section 4 names JST PH housings for J_CAM, J_QMX, J_POD and the three sensor modules and SH housings for board E's two mixer fans, and the netlists draw 2.54 mm pin header lands for all of them. Board B's ten bench and commissioning headers are owed under the same item: whether a header is fitted on them at all is the same choice)
   |   INCONCLUSIVE A: open item REL-O-07 holds the board: the expected number of mates of each connector over a service life is stated nowhere (REQ-028: no life requirement for prototype 1), so this list carries ratings and compares them with nothing (next action: when a service life is ruled, state the expected mates per connector from CONOPS section 5 and compare each class's figure with it)
   |   INCONCLUSIVE A: open item REL-O-08 holds the board: the joints under heavy soldered parts (the soldered radio modules, the magnetics, the large inductors) are joints that carry load in transport, and this inventory cannot find them: a netlist carries no mass (next action: list the parts above a mass limit from the makers' documents and add them as a class per board with the staking or support each needs)
   |   INCONCLUSIVE A: open item REL-O-13 holds the board: the inventory of a board with a schematic is its NETLIST's, and the declared-phase board files carry footprints no netlist holds: mounting holes H1 to H8 on board A, twenty on board B (M2.5, M3 and M4) with six S_ references beside them, H1 to H4 on boards D and P and twenty-eight on board E, every H on a MountingHole land, while boards C and E5 class the same kind of joint because their own artefacts carry it. The board files also carry a few R, Q, C and U references the netlists do not, and the netlists carry parts the board files do not (225 on board A), so the two are different generations of each design (next action: when each board file is regenerated from its declared netlist, read its footprints beside the netlist (wear_inventory.read_board) and class every screw joint per board with its torque, its thread lock and what hangs on it, from ASSEMBLY.md)
   |   INCONCLUSIVE A: class JST VH power headers has no cycle figure: the maker's documents that were read state none (v2/vendor/connectors/jst-vh-catalogue.pdf, v2/vendor/connectors/jst-handling-precautions-2020.pdf), so the class is undecided and the board is not passed on it (open item REL-O-12: prepare the question to each maker for the owner to send (outside contact is his), or take each class's figure from the prototype's mate-cycle test once TEST-PLAN.md sets its cycle count; carry the figure with its document, or with the test's record)
   |   INCONCLUSIVE A: class JST XH lead headers has no cycle figure: the maker's documents that were read state none (v2/vendor/connectors/jst-xh-catalogue.pdf, v2/vendor/connectors/jst-handling-precautions-2020.pdf), so the class is undecided and the board is not passed on it (open item REL-O-12: prepare the question to each maker for the owner to send (outside contact is his), or take each class's figure from the prototype's mate-cycle test once TEST-PLAN.md sets its cycle count; carry the figure with its document, or with the test's record)
   |   INCONCLUSIVE A: class JST PH lead header has no cycle figure: the maker's documents that were read state none (v2/vendor/connectors/jst-ph-catalogue.pdf, v2/vendor/connectors/jst-handling-precautions-2020.pdf), so the class is undecided and the board is not passed on it (open item REL-O-12: prepare the question to each maker for the owner to send (outside contact is his), or take each class's figure from the prototype's mate-cycle test once TEST-PLAN.md sets its cycle count; carry the figure with its document, or with the test's record)
   |   INCONCLUSIVE A: class the blade fuse holder has no cycle figure: the maker's documents that were read state none (v2/vendor/keystone/M65p42.pdf), so the class is undecided and the board is not passed on it (open item REL-O-12: prepare the question to each maker for the owner to send (outside contact is his), or take each class's figure from the prototype's mate-cycle test once TEST-PLAN.md sets its cycle count; carry the figure with its document, or with the test's record)
   | verdict: reliability            INCONCLUSIVE of 0 {"boards": 1, "candidates": 0, "citations_unjudged": 0, "classed": 0, "classes": 11, "classes_undecided": 4, "covered": 0, "excluded": 0, "exclusions": 1, "fail": 0, "figures_cited": 5, "figures_none_published": 4, "figures_not_mated": 0, "figures_owed": 2, "inconclusive": 10, "measures_owed": 0, "per_board": {"a": {"artefact": null, "bound": false, "candidates": 0, "citations_unjudged": 0, "classed": 0, "classes_undecided": 4, "excluded": 0, "held_by": ["REL-O-01", "REL-O-02", "REL-O-07", "REL-O-08", "REL-O-12", "REL-O-13"], "refused": 0, "result": "INCONCLUSIVE"}}, "refused": 0} | every candidate part of the inventory falls in one declared class, with its cycle figure from the maker's document or the reason it has none, its load and the measure taken, or under one declared exclusion with its reason. A desk reading of a netlist and a list: it tests nothing and replaces no physical verification; REL-001 is verified at the prototype and no board has been built

the matrix: 4 of 4 case(s) as wanted, 0 not

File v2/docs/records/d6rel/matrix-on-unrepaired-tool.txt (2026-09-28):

THE FOUR-CASE MATRIX ON THE UNREPAIRED TOOL (worker d6rel, MESHSAT-1357, first taken 27 September 2026 23:57 CEST, re-taken 28 September 2026 17:55 CEST with the final matrix.py)
The tool is git show 73ae2f21:v2/ecad/tools/reliability.py written to $SP/old/ ($SP is the session's scratch directory, outside the tree);
case 4's list is git show 73ae2f21:v2/ecad/tools/pcb_reliability.yaml beside it. Command, from anywhere:
  python3 v2/docs/records/d6rel/matrix.py v2/ecad/tools $SP/old/reliability.py
Exit code of the matrix script: 1 (two of the four cases are not as wanted: cases 3 and 4, the reviewer's two silent cases). The sheets are as the reviewer wrote them (no pin: the unrepaired tool knows no such key).
Nothing was built or measured: these are readings of fixture netlists.

tool under test : $SP/old/reliability.py  sha256/16 71d0872195905c9d
tools directory : <worktree>/v2/ecad/tools
case 4's list   : $SP/old/pcb_reliability.yaml  sha256/16 fbf56eb06df1d007
fixtures in     : a temporary directory outside the tree (mkdtemp prefix d6rel-matrix-)

== case 1-one-declared-jst: one declared JST connector
   wanted PASS (exit 0); the tool says PASS (exit 0): as wanted
   counts {"boards": 1, "classes": 1, "covered": 1, "fail": 0}  denominator 2  missing_input None
   inputs recorded: {"board": "a", "list": {"path": "list.yaml", "sha256_16": "fa012ad00726698c"}}
   | reliability: A    1 class(es),  1 part(s) covered
   | verdict: reliability            PASS         of 2 {"boards": 1, "classes": 1, "covered": 1, "fail": 0} | every part that carries load or sees cycling falls in a declared class with its cycle figure or the reason it has none, its load and the measure taken. It tests nothing: REL-001 is verified at the prototype and no board has been built

== case 2-plus-undeclared-idc: plus an undeclared IDC header
   wanted FAIL (exit 1); the tool says FAIL (exit 1): as wanted
   counts {"boards": 1, "classes": 1, "covered": 1, "fail": 1}  denominator 2  missing_input None
   inputs recorded: {"board": "a", "list": {"path": "list.yaml", "sha256_16": "fa012ad00726698c"}}
   | reliability: A    1 class(es),  1 part(s) covered
   |   FAIL A: J_RIB1 (fixture ribbon (IDC 2x5)) carries load or sees cycling and is in no declared class
   | verdict: reliability            FAIL         of 2 {"boards": 1, "classes": 1, "covered": 1, "fail": 1} | every part that carries load or sees cycling falls in a declared class with its cycle figure or the reason it has none, its load and the measure taken. It tests nothing: REL-001 is verified at the prototype and no board has been built

== case 3-plus-undeclared-rj45: plus an undeclared "RJ45 MagJack"
   wanted FAIL (exit 1); the tool says PASS (exit 0): NOT AS WANTED
   counts {"boards": 1, "classes": 1, "covered": 1, "fail": 0}  denominator 2  missing_input None
   inputs recorded: {"board": "a", "list": {"path": "list.yaml", "sha256_16": "fa012ad00726698c"}}
   | reliability: A    1 class(es),  1 part(s) covered
   | verdict: reliability            PASS         of 2 {"boards": 1, "classes": 1, "covered": 1, "fail": 0} | every part that carries load or sees cycling falls in a declared class with its cycle figure or the reason it has none, its load and the measure taken. It tests nothing: REL-001 is verified at the prototype and no board has been built

== case 4-board-a-no-netlist: board A's declaration and no netlist
   wanted INCONCLUSIVE (exit 3); the tool says PASS (exit 0): NOT AS WANTED
   counts {"boards": 1, "classes": 6, "covered": 0, "fail": 0}  denominator 6  missing_input None
   inputs recorded: {"board": "a", "list": {"path": "list.yaml", "sha256_16": "fbf56eb06df1d007"}}
   | reliability: A    6 class(es),  0 part(s) covered  (no netlist here)
   |   note board A has no netlist in this tree, so the list could not be compared with it
   | verdict: reliability            PASS         of 6 {"boards": 1, "classes": 6, "covered": 0, "fail": 0} | every part that carries load or sees cycling falls in a declared class with its cycle figure or the reason it has none, its load and the measure taken. It tests nothing: REL-001 is verified at the prototype and no board has been built

the matrix: 2 of 4 case(s) as wanted, 2 not

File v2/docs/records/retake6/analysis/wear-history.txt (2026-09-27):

retake6: why boards D, E and P each count one more covered part than their readings of 21 September 2026 (written by wear_history.py, read only)
The readings of 21 September: D 9 (12:51:26Z), E 7 (12:52:10Z), P 6 (12:52:46Z). The re-take: D 10, E 8, P 7.

8ce0b892  v2/ecad/pcb-d-aprs-d9/out/pcb-d-aprs.net: wear set 9, covered by exactly one declared class 9, classes declared 3 (the radio module's sockets; the antenna jack and the PA ports; the power and harness headers)
824ec9d4  v2/ecad/pcb-d-aprs-d9/out/pcb-d-aprs.net: wear set 9, covered by exactly one declared class 9, classes declared 3 (the radio module's sockets; the antenna jack and the PA ports; the power and harness headers)
232231be  v2/ecad/pcb-d-aprs-d9/out/pcb-d-aprs.net: wear set 9, covered by exactly one declared class 9, classes declared 3 (the radio module's sockets; the antenna jack and the PA ports; the power and harness headers)
faf8c981  v2/ecad/pcb-d-aprs-d9/out/pcb-d-aprs.net: wear set 9, covered by exactly one declared class 9, classes declared 3 (the radio module's sockets; the antenna jack and the PA ports; the power and harness headers)
458b2873  v2/ecad/pcb-d-aprs-d9/out/pcb-d-aprs.net: wear set 9, covered by exactly one declared class 9, classes declared 3 (the radio module's sockets; the antenna jack and the PA ports; the power and harness headers)
76235aad  v2/ecad/pcb-d-aprs-d9/out/pcb-d-aprs.net: wear set 10, covered by exactly one declared class 10, classes declared 4 (the radio module's sockets; the antenna jack and the PA ports; the power and harness headers; the power amplifier's flange NTC lead)
     + J_FLANGE   JST-XH 1x2 socket: power amplifier flange NTC lead (Semitec 103AT-2 on the flange, bench-fitted): NTC GND
b7f96784  v2/ecad/pcb-d-aprs-d9/out/pcb-d-aprs.net: wear set 10, covered by exactly one declared class 10, classes declared 4 (the radio module's sockets; the antenna jack and the PA ports; the power and harness headers; the power amplifier's flange NTC lead)
6ec37197  v2/ecad/pcb-d-aprs-d9/out/pcb-d-aprs.net: wear set 10, covered by exactly one declared class 10, classes declared 4 (the radio module's sockets; the antenna jack and the PA ports; the power and harness headers; the power amplifier's flange NTC lead)
73ae2f21  v2/ecad/pcb-d-aprs-d9/out/pcb-d-aprs.net: wear set 10, covered by exactly one declared class 10, classes declared 4 (the radio module's sockets; the antenna jack and the PA ports; the power and harness headers; the power amplifier's flange NTC lead)

d58b8d45  v2/ecad/pcb-e1-dock-e7/out/pcb-e1-dock.net: wear set 7, covered by exactly one declared class 7, classes declared 3 (the pack lead connector; the blade fuse holders; the DC inlet, the solar input and the SMBus header)
824ec9d4  v2/ecad/pcb-e1-dock-e7/out/pcb-e1-dock.net: wear set 7, covered by exactly one declared class 7, classes declared 3 (the pack lead connector; the blade fuse holders; the DC inlet, the solar input and the SMBus header)
faf8c981  v2/ecad/pcb-e1-dock-e7/out/pcb-e1-dock.net: wear set 8, covered by exactly one declared class 8, classes declared 3 (the pack lead connector; the blade fuse holders; the DC inlet, the solar input, the SMBus header and the lid sensor lead)
     + J_TAMP     JST-XH 1x2 (B2B-XH-A): lid and tamper reed sensor lead, Littelfuse 59140-1-S-05-A normally open under the frame, 57140-000 magnet in the lid: 1 lead, 
bc0f562f  v2/ecad/pcb-e1-dock-e7/out/pcb-e1-dock.net: wear set 8, covered by exactly one declared class 8, classes declared 3 (the pack lead connector; the blade fuse holders; the DC inlet, the solar input, the SMBus header and the lid sensor lead)
b7f96784  v2/ecad/pcb-e1-dock-e7/out/pcb-e1-dock.net: wear set 8, covered by exactly one declared class 8, classes declared 3 (the pack lead connector; the blade fuse holders; the DC inlet, the solar input, the SMBus header and the lid sensor lead)
6ec37197  v2/ecad/pcb-e1-dock-e7/out/pcb-e1-dock.net: wear set 8, covered by exactly one declared class 8, classes declared 3 (the pack lead connector; the blade fuse holders; the DC inlet, the solar input, the SMBus header and the lid sensor lead)
73ae2f21  v2/ecad/pcb-e1-dock-e7/out/pcb-e1-dock.net: wear set 8, covered by exactly one declared class 8, classes declared 3 (the pack lead connector; the blade fuse holders; the DC inlet, the solar input, the SMBus header and the lid sensor lead)

a0b707f9  v2/ecad/pcb-p-pack-p2/out/pcb-p-pack.net: wear set 6, covered by exactly one declared class 6, classes declared 3 (the pack terminals; the cell tap and thermistor headers; the pack fuse holder)
faf8c981  v2/ecad/pcb-p-pack-p2/out/pcb-p-pack.net: wear set 6, covered by exactly one declared class 6, classes declared 3 (the pack terminals; the cell tap and thermistor headers; the pack fuse holder)
d90f30e4  v2/ecad/pcb-p-pack-p2/out/pcb-p-pack.net: wear set 7, covered by exactly one declared class 7, classes declared 3 (the pack terminals; the cell tap and thermistor headers; the pack fuse holder)
     + J_TS2      second-level cell thermistor socket, JST-PH 1x2 (Semitec 103AT-2 on the hottest cell): 1 TS_SEC_J, 2 VSS
7bef62bd  v2/ecad/pcb-p-pack-p2/out/pcb-p-pack.net: wear set 7, covered by exactly one declared class 7, classes declared 3 (the pack terminals; the cell tap and thermistor headers; the pack fuse holder)
6ec37197  v2/ecad/pcb-p-pack-p2/out/pcb-p-pack.net: wear set 7, covered by exactly one declared class 7, classes declared 3 (the pack terminals; the cell tap and thermistor headers; the pack fuse holder)
73ae2f21  v2/ecad/pcb-p-pack-p2/out/pcb-p-pack.net: wear set 7, covered by exactly one declared class 7, classes declared 3 (the pack terminals; the cell tap and thermistor headers; the pack fuse holder)

6ec37197  v2/ecad/pcb-b-compute-b19/out/pcb-b-compute.net: wear set 38, covered by exactly one declared class 38, classes declared 6 (CM5 module receptacles; M.2 sockets; U.FL antenna sockets; the coin cell holder; fan and flash headers, the panel ribbon, the HDMI and USB receptacles; the PCIe switches' own sockets on the carrier)
73ae2f21  v2/ecad/pcb-b-compute-b19/out/pcb-b-compute.net: wear set 38, covered by exactly one declared class 38, classes declared 6 (CM5 module receptacles; M.2 sockets; U.FL antenna sockets; the coin cell holder; fan and flash headers, the panel ribbon, the HDMI and USB receptacles; the PCIe switches' own sockets on the carrier)

6ec37197  v2/ecad/pcb-a-power-a23/out/pcb-a-power.net: wear set 39, covered by exactly one declared class 39, classes declared 6 (SMA bulkhead jacks; blind-mate dock contacts; JST-VH power headers; IDC ribbon headers; the main switch and USB-C wall leads; the blade fuse holder)
73ae2f21  v2/ecad/pcb-a-power-a23/out/pcb-a-power.net: wear set 39, covered by exactly one declared class 39, classes declared 6 (SMA bulkhead jacks; blind-mate dock contacts; JST-VH power headers; IDC ribbon headers; the main switch and USB-C wall leads; the blade fuse holder)
6ec37197  v2/ecad/pcb-c-display-c8/out/pcb-c-display.net: wear set 9, covered by exactly one declared class 9, classes declared 2 (the panel ribbon header; the face plate's mounting holes)
73ae2f21  v2/ecad/pcb-c-display-c8/out/pcb-c-display.net: wear set 9, covered by exactly one declared class 9, classes declared 2 (the panel ribbon header; the face plate's mounting holes)

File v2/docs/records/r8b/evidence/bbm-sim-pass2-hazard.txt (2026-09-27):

requirement: lead >= 1.000 us, hold >= 40.000 us
netlist BOX/out/t8/regen/pcb-b-compute.net: 46 gates, 12 Schmitt buffers, 9 RC nodes; hazard model ON
  1 single vote change (corners)                   runs   162  select moves    162  min lead 426.896 us  min hold 392.802 us  violations 0
  2 vote returns after r (checker's case)          runs 17009  select moves  50564  min lead 249.422 us  min hold 194.464 us  violations 0
  3 adversary aimed at the circuit's instants      runs   450  select moves   1344  min lead 46.505 us  min hold 227.008 us  violations 0
  4 random vote waveforms                          runs  3181  select moves   8344  min lead 73.226 us  min hold 249.405 us  violations 0
  4 random vote waveforms with power-good toggles  runs  1319  select moves   3366  min lead 82.147 us  min hold 332.419 us  violations 0
TOTAL runs 22121, select moves 63780, violations 0

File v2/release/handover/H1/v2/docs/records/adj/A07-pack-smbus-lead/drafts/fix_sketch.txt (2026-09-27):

A07 minimum fix sketch (not applied; one writer per file, condition 4; each regeneration proven by a netlist diff, condition 5)
E (gen_sch_e.py):
  :117-120 FP.update add  "XH4": "Connector_JST:JST_XH_B4B-XH-A_1x04_P2.50mm_Vertical"
  :136 replace ph("J_SMB", 6, ...) with
       part("J_SMB", "Connector_Generic", "Conn_01x04", "SMBus lead from P1 J_SMB (JST-XH 1x4): SCL0 SDA0 GND, pin 4 PRES not connected", "XH4", {"1": "SCL0", "2": "SDA0", "3": "GND", "4": "NC"})
       (lcsc_fill.py:158 then assigns C594232 by re.match on the value and JST_XH_B4B in the footprint, lcsc_fill.py:238)
  pcb-e1-dock*/lcsc-allow.txt:7 "(XH or pin header)" line removed
  :131 and :349 comments: no BB-2590 sections; GPIO2/3 are the RP2040's I2C1 block, GPIO4/5 its I2C0 (Table 279)
  parity: netlist diff shows only J_SMB (footprint, pins 1 and 2 swapped roles onto SCL0/SDA0, SDA1/SCL1 lose J_SMB, one GND pin)
P (gen_sch_p.py):
  :172 J_SMB pin 3 GND -> PACK_N (TI SLUSC67B Figure 21: J2 VSS on CHGND with J4 PACK-, not the cell-side GND)
  :171 D2 (separate defect, own issue): VBUS pin 5 is on VCC_F (PACK_P through R7 1k, 12 to 16.8 V) against USBLC6-2 VRM 5.25 V / VBR 6 V;
       TI's own arrangement is two 5.6 V zeners (MM3Z5V6C) from SMBC and SMBD to the pack-side ground (Figures 21 and 30)
  parity: netlist diff shows only J_SMB.3 (and D2 if taken)
Lead: JST XH 1x4 at both ends, pin n to pin n, 26 AWG twisted, 350 mm
Docs: ASSEMBLY.md:45, :60, :140; PANEL.md:128, :155; a new appendix entry correcting 32.62 (line 3062) rather than editing it
Gate: check_contracts.py gets a J_SMB contract (today 0 occurrences): same family, pitch, count, and pin n role equal on P and E

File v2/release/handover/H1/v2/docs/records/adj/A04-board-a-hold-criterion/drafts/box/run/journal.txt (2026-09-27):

A04 journal 2026-09-25T21:30:08Z host d7e94791178c clone 82dd1e4dc44efabeee1164a995cda4e866610f3d main-clone 82dd1e4dc44efabeee1164a995cda4e866610f3d
== 1. part-for-part comparison
A04 part-for-part comparison, board A, commit 82dd1e4dc44efabeee1164a995cda4e866610f3d, pcbnew 9.0.9
  netlist     v2/ecad/pcb-a-power-a23/out/pcb-a-power.net sha256 aa1372ba3932610f (worktree aa1372ba3932610f) last 0d1e2ef6 2026-09-20T14:23:13+02:00
  board       v2/ecad/pcb-a-power-a23/pcb-a-power.kicad_pcb sha256 58e26c67987b1daa (worktree 58e26c67987b1daa) last b7e0d28f 2026-09-15T07:50:52+02:00
  intent      v2/ecad/pcb-a-power-a23/out/pcb-a-power-intent.json sha256 abeb227d673b3af3 (worktree abeb227d673b3af3) last 0d1e2ef6 2026-09-20T14:23:13+02:00
  board_table v2/ecad/tools/boards/a.json sha256 0fd6672749bc8875 (worktree 0fd6672749bc8875) last 1bf7fca1 2026-09-21T23:45:42+02:00
  board phase texts: ['MESHSAT FIELD KIT  -  PCB-A POWER + I/O  -  REV A (A32)'] ; boards/a.json phase A32
conductors: J_DOCK.1=VIN_RAW, J_DOCK.2=VIN_RAW, J_DOCK.3=VIN_RAW(same net, undeclared pin), J_DOCK.4=VIN_RAW(same net, undeclared pin), J_USBW.1=USB_WALL_P, J_USBW.2=USB_WALL_N, J_USBC_OUT.1=PD_VBUS, J_USBC_OUT.2=PD_CC1, J_USBC_OUT.3=PD_CC2

ref         verdict    role      | netlist value || board value | footprint nl / board | land | pad nets
C11         DIFFERENT  on the conductor           | 10u 100V X7R 1210 || 10u 50V X7R 1210 | Capacitor_SMD:C_1210_3225Metric / C_1210_3225Metric | IDENTICAL to Capacitor_SMD:C_1210_3225Me | all 2 equal
            lcsc netlist None board None; board F.Cu at (35.0, 45.5) rot 90.0
C12         DIFFERENT  on the conductor           | 10u 100V X7R 1210 || 10u 50V X7R 1210 | Capacitor_SMD:C_1210_3225Metric / C_1210_3225Metric | IDENTICAL to Capacitor_SMD:C_1210_3225Me | all 2 equal
            lcsc netlist None board None; board F.Cu at (35.0, 51.0) rot 90.0
C120        SAME       on the conductor           | 10u 25V 1210 || 10u 25V 1210 | Capacitor_SMD:C_1210_3225Metric / C_1210_3225Metric | IDENTICAL to Capacitor_SMD:C_1210_3225Me | all 2 equal
            lcsc netlist None board None; board F.Cu at (161.835, 56.975) rot 0.0
C96         SAME       on the conductor           | 330p || 330p | Capacitor_SMD:C_0603_1608Metric / C_0603_1608Metric | IDENTICAL to Capacitor_SMD:C_0603_1608Me | all 2 equal
            lcsc netlist None board None; board F.Cu at (152.105, 61.215) rot 0.0
C97         SAME       on the conductor           | 330p || 330p | Capacitor_SMD:C_0603_1608Metric / C_0603_1608Metric | IDENTICAL to Capacitor_SMD:C_0603_1608Me | all 2 equal
            lcsc netlist None board None; board F.Cu at (156.315, 61.215) rot 0.0
D2          DIFFERENT  PROTECTION                 | SMCJ40A (VIN_RAW clamp behind E6's filter: 40 V standoff on a line spe || SMCJ33A (VIN_RAW clamp behind E6's filter) | Diode_SMD:D_SMC / D_SMC | IDENTICAL to Diode_SMD:D_SMC | all 2 equal
            polarity: {"perpendicular_silk_offsets_toward_pad1_mm": [4.91], "cathode_mark_beside": "pad 1", "netlist_pad1": "VIN_RAW", "netlist_pad2": "GND", "board_pad1": ["VIN_RAW"], "board_pad2": ["GND"], "library_cathode_mark_beside": "pad 1"}
            lcsc netlist C224052 board None; board F.Cu at (37.57, 69.475) rot 0.0
D4          SAME       PROTECTION                 | SMBJ18A (VBUS clamp at the outlet) || SMBJ18A (VBUS clamp at the outlet) | Diode_SMD:D_SMB / D_SMB | IDENTICAL to Diode_SMD:D_SMB | all 2 equal
            polarity: {"perpendicular_silk_offsets_toward_pad1_mm": [3.66], "cathode_mark_beside": "pad 1", "netlist_pad1": "PD_VBUS", "netlist_pad2": "GND", "board_pad1": ["PD_VBUS"], "board_pad2": ["GND"], "library_cathode_mark_beside": "pad 1"}
            lcsc netlist None board None; board F.Cu at (163.06, 50.875) rot 0.0
J_AB2       SAME       on the conductor           | A-B wall-port ribbon (IDC 2x5): the wall USB pair on the END row with  || A-B wall-port ribbon (IDC 2x5): the wall USB pair on the END row with  | meshsat:IDC-Header_2x05_P2.54mm_Vertical_NarrowPad / IDC-Header_2x05_P2.54mm_Vertical_NarrowPad | IDENTICAL to meshsat:IDC-Header_2x05_P2. | all 10 equal
            lcsc netlist None board None; board F.Cu at (245.752, 126.08) rot 180.0
J_DOCK      SAME       port connector             | spring pins to the dock block (2x6, Preci-Dip 813-S1-012-10-016101, un || spring pins to the dock block (2x6, Preci-Dip 813-S1-012-10-016101, un | meshsat:PogoPins_2x6 / PogoPins_2x6 | IDENTICAL to meshsat:PogoPins_2x6 | all 12 equal
            lcsc netlist None board None; board B.Cu at (74.0, 180.0) rot 0.0
J_USBC_OUT  SAME       port connector             | wall USB-C outlet, power side (pigtail header): VBUS CC1 CC2 GND GND || wall USB-C outlet, power side (pigtail header): VBUS CC1 CC2 GND GND | Connector_PinHeader_2.54mm:PinHeader_1x05_P2.54mm_Vertical / PinHeader_1x05_P2.54mm_Vertical | IDENTICAL to Connector_PinHeader_2.54mm: | all 5 equal
            lcsc netlist None board None; board F.Cu at (254.92, 84.0) rot 90.0
J_USBW      SAME       port connector             | JST-PH 1x4 socket: the wall USB-C data pair to B16 passes here on the  || JST-PH 1x4 socket: the wall USB-C data pair to B16 passes here on the  | Connector_JST:JST_PH_B4B-PH-K_1x04_P2.00mm_Vertical / JST_PH_B4B-PH-K_1x04_P2.00mm_Vertical | IDENTICAL to Connector_JST:JST_PH_B4B-PH | all 4 equal
            lcsc netlist C131334 board None; board F.Cu at (259.45, 125.0) rot 90.0
Q2          SAME       on the conductor           | CSD19532Q5B 100 V N-FET (4.6 mOhm at VGS 6 V, PowerPAK SO-8 / SON-8 5x || CSD19532Q5B 100 V N-FET (4.6 mOhm at VGS 6 V, PowerPAK SO-8 / SON-8 5x | Package_SO:PowerPAK_SO-8_Single / PowerPAK_SO-8_Single | IDENTICAL to Package_SO:PowerPAK_SO-8_Si | all 5 equal
            lcsc netlist C473333 board None; board F.Cu at (42.195, 45.5) rot 0.0
R138        SAME       on the conductor           | 10mOhm 1% 2512 (ISNS) || 10mOhm 1% 2512 (ISNS) | Resistor_SMD:R_2512_6332Metric / R_2512_6332Metric | IDENTICAL to Resistor_SMD:R_2512_6332Met | all 2 equal
            lcsc netlist None board None; board F.Cu at (171.79, 50.555) rot 0.0
R139        SAME       on the conductor           | 43R 1W 2512 (DSCG) || 43R 1W 2512 (DSCG) | Resistor_SMD:R_2512_6332Metric / R_2512_6332Metric | IDENTICAL to Resistor_SMD:R_2512_6332Met | all 2 equal
            lcsc netlist None board None; board F.Cu at (154.455, 57.305) rot 0.0
R14         SAME       on the conductor           | 62k 1% || 62k 1% | Resistor_SMD:R_0603_1608Metric / R_0603_1608Metric | IDENTICAL to Resistor_SMD:R_0603_1608Met | all 2 equal
            lcsc netlist None board None; board F.Cu at (38.315, 78.555) rot 0.0
TP13        SAME       on the conductor           | VIN_RAW || VIN_RAW | TestPoint:TestPoint_Pad_D1.5mm / TestPoint_Pad_D1.5mm | IDENTICAL to TestPoint:TestPoint_Pad_D1. | all 1 equal
            lcsc netlist None board None; board F.Cu at (37.625, 75.325) rot 0.0
U18         SAME       protection inside part (decision 31 declaration) | TPS25740ARGER USB-C PD source controller, 45 W outlet (5, 9, 15 V at 3 || TPS25740ARGER USB-C PD source controller, 45 W outlet (5, 9, 15 V at 3 | Package_DFN_QFN:QFN-24-1EP_4x4mm_P0.5mm_EP2.5x2.5mm / QFN-24-1EP_4x4mm_P0.5mm_EP2.5x2.5mm | IDENTICAL to Package_DFN_QFN:QFN-24-1EP_ | all 25 equal
            lcsc netlist C544309 board None; board F.Cu at (160.188, 45.0) rot 0.0
U2          DIFFERENT  on the conductor           | LM5176PWPR buck-boost controller, VBUS20 from VIN_RAW || LM5176PWPR buck-boost controller, VBUS20 from VIN_RAW | Package_SO:HTSSOP-28-1EP_4.4x9.7mm_P0.65mm_EP2.85x5.4mm / HTSSOP-28-1EP_4.4x9.7mm_P0.65mm_EP2.85x5.4mm | IDENTICAL to Package_SO:HTSSOP-28-1EP_4. | pin 13: netlist FE_ISNS_N, board ['VBUS20']; pin 14: netlist FE_ISNS_P, board ['FE_OUT']; pin 15: netlist FE_CSGF, board ['GND']; pin 16: netlist FE_CSF, board ['FE_CS']
            lcsc netlist C442493 board None; board F.Cu at (56.0, 54.047) rot 0.0
U29         SAME       PROTECTION                 | USBLC6-2SC6 || USBLC6-2SC6 | Package_TO_SOT_SMD:SOT-23-6 / SOT-23-6 | IDENTICAL to Package_TO_SOT_SMD:SOT-23-6 | all 6 equal
            lcsc netlist C7519 board None; board F.Cu at (253.088, 125.0) rot 90.0

net PD_CC1      equal=True netlist_only=[] board_only=[] nodes=['C96.1', 'J_USBC_OUT.2', 'U18.2']
net PD_CC2      equal=True netlist_only=[] board_only=[] nodes=['C97.1', 'J_USBC_OUT.3', 'U18.3']
net PD_VBUS     equal=True netlist_only=[] board_only=[] nodes=['C120.1', 'D4.1', 'J_USBC_OUT.1', 'R138.2', 'R139.2', 'U18.21']
net USB_WALL_N  equal=True netlist_only=[] board_only=[] nodes=['J_AB2.2', 'J_USBW.2', 'U29.3', 'U29.4']
net USB_WALL_P  equal=True netlist_only=[] board_only=[] nodes=['J_AB2.1', 'J_USBW.1', 'U29.1', 'U29.6']
net VIN_RAW     equal=True netlist_only=[] board_only=[] nodes=['C11.1', 'C12.1', 'D2.1', 'J_DOCK.1', 'J_DOCK.2', 'J_DOCK.3', 'J_DOCK.4', 'Q2.5', 'R14.1', 'TP13.1', 'U2.2', 'U2.3']

TRN-001 walk on committed netlist: fail=[] in_part=2
TRN-001 walk on the BOARD's own connectivity and values: fail=[] in_part=2
values swapped into board-values netlist: 3, e.g. ['C11', 'C12', 'D2']
exit 0
== 2. TRN-001 fresh on the committed netlist (port_protect.py)
port_protect: board A declares 3 external port(s); 3 found on this netlist
  J_DOCK       12 pin(s), 0 unprotected, 0 behind an active part, 0 answered in the part it reaches  [shore and vehicle DC arriving over the dock from the wall recept]
  J_USBW       4 pin(s), 0 unprotected, 0 behind an active part, 0 answered in the part it reaches  [the wall USB host port through the MIL-DTL-38999 receptacle: a p]
  J_USBC_OUT   5 pin(s), 0 unprotected, 0 behind an active part, 2 answered in the part it reaches  [the USB-C outlet on the connector plate, out of the case]
      ANSWERED J_USBC_OUT.2 on PD_CC1: protection inside U18, cited: TI TPS25740A datasheet, v2/vendor/ti/ti-tps25740.pdf section 9.1.1 System-Level ESD Protection: 'The device has ESD protection built into the CC1 and CC2 pins so that no external protection is necessary.' Its absolute maximum on CC1 and CC2 is -0.3 to 6 V, and the VBUS path its own Figure 37 clamps is D4, an SMBJ18A, which this board already carries. Owner decision 31, ruled by the session on 21 September 2026 against the IEC 61000-4-2 level 4 that decision 34 states.
      ANSWERED J_USBC_OUT.3 on PD_CC2: protection inside U18, cited: TI TPS25740A datasheet, v2/vendor/ti/ti-tps25740.pdf section 9.1.1 System-Level ESD Protection: 'The device has ESD protection built into the CC1 and CC2 pins so that no external protection is necessary.' Its absolute maximum on CC1 and CC2 is -0.3 to 6 V, and the VBUS path its own Figure 37 clamps is D4, an SMBJ18A, which this board already carries. Owner decision 31, ruled by the session on 21 September 2026 against the IEC 61000-4-2 level 4 that decision 34 states.
verdict: port_protect           PASS         of 21 {"answered_in_part": 2, "behind_an_active_part": 0, "declared": 3, "not_on_netlist": 0, "ports": 3, "unprotected": 0} | every declared external conductor meets a protection part before a chip
exit 0
== 3. SCH-002 fresh: committed board against committed netlist (netlist_board.py)
netlist_board: FAIL C121 is in the netlist and not on the board
netlist_board: FAIL C122 is in the netlist and not on the board
netlist_board: FAIL C123 is in the netlist and not on the board
netlist_board: FAIL C124 is in the netlist and not on the board
netlist_board: FAIL C125 is in the netlist and not on the board
netlist_board: FAIL C126 is in the netlist and not on the board
netlist_board: FAIL C127 is in the netlist and not on the board
netlist_board: FAIL C128 is in the netlist and not on the board
netlist_board: FAIL C129 is in the netlist and not on the board
netlist_board: FAIL C130 is in the netlist and not on the board
netlist_board: FAIL C131 is in the netlist and not on the board
netlist_board: FAIL C132 is in the netlist and not on the board
netlist_board: FAIL R146 is in the netlist and not on the board
netlist_board: FAIL R147 is in the netlist and not on the board
netlist_board: FAIL R148 is in the netlist and not on the board
netlist_board: FAIL R149 is in the netlist and not on the board
netlist_board: FAIL R150 is in the netlist and not on the board
netlist_board: FAIL R151 is in the netlist and not on the board
netlist_board: FAIL R152 is in the netlist and not on the board
netlist_board: FAIL R153 is in the netlist and not on the board
netlist_board: FAIL R154 is in the netlist and not on the board
netlist_board: FAIL R155 is in the netlist and not on the board
netlist_board: FAIL R156 is in the netlist and not on the board
netlist_board: FAIL R157 is in the netlist and not on the board
netlist_board: FAIL R158 is in the netlist and not on the board
netlist_board: FAIL R159 is in the netlist and not on the board
netlist_board: FAIL R160 is in the netlist and not on the board
netlist_board: FAIL R161 is in the netlist and not on the board
netlist_board: FAIL R162 is in the netlist and not on the board
netlist_board: FAIL R163 is in the netlist and not on the board
netlist_board: 1980 of 2040 comparisons agree (428 references in the netlist, 400 footprints on the board)
verdict: netlist_board          FAIL         of 2040 {"agree": 1980, "aliased_pins": 0, "board_footprints": 400, "board_only_inert": 0, "fail": 60, "netlist_refs": 428} | the board against the schematic it was placed from
exit 1
== 4. CMP-001 on the committed netlist (derate.py)
derate: 144 rated part-on-net pair(s) judged at a 20% margin over 27 declared rail(s) and 52 declared node(s), 0 of them against the part maker's own reference circuit; 77 part(s) carry no rating in their value and were not judged; 0 net(s) carry a rated part and no declared voltage
verdict: derate                 PASS         of 144 {"by_vendor_reference": 0, "judged": 144, "undeclared_nets": 0, "under_rated": 0, "unrated_parts": 77} | a part's rating against the declared voltage of the rail it is soldered to; DC-bias capacitance derating is NOT checked here and is an open gap
exit 0
== 5. CMP-001 on the same netlist carrying the BOARD's values (derate.py)
derate: 144 rated part-on-net pair(s) judged at a 20% margin over 27 declared rail(s) and 52 declared node(s), 0 of them against the part maker's own reference circuit; 77 part(s) carry no rating in their value and were not judged; 0 net(s) carry a rated part and no declared voltage
  FAIL D2 (SMCJ33A (VIN_RAW clamp behind E6's filter)) stands off 33.0 V and protects VIN_RAW, which runs to 36.0 V in normal service: it conducts in service rather than only on a transient
verdict: derate                 FAIL         of 144 {"by_vendor_reference": 0, "judged": 144, "undeclared_nets": 0, "under_rated": 1, "unrated_parts": 77} | a part's rating against the declared voltage of the rail it is soldered to; DC-bias capacitance derating is NOT checked here and is an open gap
exit 1
== 6. the clone is untouched
done 2026-09-25T21:30:15Z

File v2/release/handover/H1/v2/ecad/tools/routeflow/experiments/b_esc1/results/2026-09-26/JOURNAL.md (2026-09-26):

# Q-B-ESC-1 journal (EXPERIMENTAL)

Board B escape trial, v2/docs/B-FEASIBILITY.md section 7. EXPERIMENTAL: never a phase, a promotion or a layout candidate.

- start: 2026-09-26T18:48:19+00:00
- commit: 44cfa0450c74e26e7e8d48261d9f7209404ccd98; tools tree: ee1906fab4cbaad78133316d1f06176288e1d8d0
- trial scripts sha256/16: run.sh a7e32b812e5b559a; count_open.py 093839e72286f50c; judge.py 0d849b2577171e79; make_arm8.py e1482746504485a7; plateau_watch.py 0a7d15af2178078e; 
- run.sh tracked at this commit: yes
- jar: freerouting-1.9.0-mesh.jar sha256/16 82753043cb9da3ae; java: openjdk version "25.0.4.1" 2026-08-18
- kicad-cli: 9.0.9; host: d7e94791178c; cores: 64
- caps: passes 20, job timeout 9000 s, first pass 5400 s, plateau 3, budget 6 h / 10 USD at 0.142 USD/h, cap 21600 s, route deadline 2026-09-27T00:03:19+00:00
- one job per arm: the router is deterministic (tests/test_driver_hygiene.py), so a repeat is the same number twice

- input: pcb-b-compute-b19/routed/pcb-b-compute-preroute.kicad_pcb sha256 62facf0952ff4c01cb0a47698ec6870b5fae0f0d9b836bf95db6c3c7bae166dd; project file sha256 c2c6e771722d9f53
make_arm8: a8 enabled copper F.Cu In1.Cu In2.Cu In3.Cu In4.Cu In5.Cu In6.Cu B.Cu; arms agree
- ESCAPE_SKIP (tools/boards/b.json escape_env): U3,U4,J_HDMI
- integrity: groups {'S1': 158, 'S2': 157, 'DEVW': 116, 'S3': 146, 'GLOBAL': 183, 'DEVE': 84} place_audit {'collisions': 10, 'fine_pitch': 75, 'footprints': 957, 'measured': 75}
- a6 pass 0: count_open: group S3 open 290 over 146 nets (135 split by the walk), residue {'U301': 36, 'U302': 8, 'U309': 5, 'U32B': 11}, vias 184, 19.9 s
- a8 pass 0: count_open: group S3 open 290 over 146 nets (135 split by the walk), residue {'U301': 36, 'U302': 8, 'U309': 5, 'U32B': 11}, vias 184, 19.9 s
- a6: route_part pid 746586 on F.Cu In2.Cu In3.Cu B.Cu, watcher pid 746587, start 2026-09-26T18:50:31+00:00
- a8: route_part pid 746595 on F.Cu In2.Cu In3.Cu In5.Cu In6.Cu B.Cu, watcher pid 746596, start 2026-09-26T18:50:31+00:00
- operator 2026-09-26T19:47:02+00:00: both routers idle since 18:50:37 on Freerouting's modal "DSN file reader" warning (net normalization); fr_watch never fired because the idle JVM's CPU ticks still move; Return sent to each display by hand, the action fr_watch is written to take
- operator watcher 2026-09-26T21:20:45+00:00: no router left, exiting
- a6: plateau_watch: stop JOB_ENDED after 12 session(s), counts [138, 111, 84, 71, 66, 56, 42, 39, 40, 37, 38, 33]
- a8: plateau_watch: stop PLATEAU after 14 session(s), counts [106, 66, 40, 28, 29, 28, 22, 25, 21, 18, 16, 23, 18, 18]
- a6 final: count_open: group S3 open 33 over 146 nets (23 split by the walk), residue {'U301': 3, 'U302': 1, 'U309': 1, 'U32B': 2}, vias 440, 8.2 s
- a6 hard set: 0 499 (H U, board-wide U includes every group the trial did not route)
- a8 final: count_open: group S3 open 18 over 146 nets (16 split by the walk), residue {'U301': 4, 'U309': 1}, vias 398, 5.8 s
- a8 hard set: 0 499 (H U, board-wide U includes every group the trial did not route)
judge: INCONCLUSIVE: an arm is not settled: it ended or was cut by a cap while its count was still falling (a6 stop JOB_ENDED, falling True; a8 stop PLATEAU, falling False)
- end: 2026-09-26T21:21:46+00:00; wall 9207 s
- fetch, file by file, then destroy the box and read the instance list: JOURNAL.md integrity.json arm8.json outcome.json and, per arm, base.json final.json s3-counts.txt s3-drc.json place_audit.txt route.log watch.log watch/passes.csv watch/watch.json run/S3/fr.log

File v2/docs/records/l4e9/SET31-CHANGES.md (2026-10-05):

**DONE:** section 8 (blocks 8 and 8a to 8g) and PC-01 to PC-16 applied to the page, the register, the generator's data and renderers, its output (regenerated through `_bin/regen_out.py`) and `test_l4e9.py`'s expectations; the overlaps reconciled to the narrower claim; `run.py test_l4e9. test_public_hygiene.` 68 passed, 0 failed, 0 skipped. **NOT DONE:** the re-pins owed at the freeze (records l4e10 and l4e11 pin this page, l6r2 the register; L4-E9's three l8p copies, PC-04), LH-12 (not this record's file), the 45.88 K/W statements outside PC-05's scope (list C). **NEXT:** the coordinator integrates after commit 2b (the cascade outputs this branch's output pins) and re-pins at the freeze.

# Set 31: L4-E9's page, register and generator brought to the set 30 candidate (MESHSAT-1357, 6 October 2026)

**Base.** `fnd/l4e9s31` from `bbba3e53e396d3fe0f8ddd2f38d0c169bcc99c45` (set 30's integration 2a on `fnd/p0pwr`: the generator re-pinned,
its D-10/D-16 citation check reading L4-E7's P0 output too). **Inputs** (read with `git show`, not in this branch): the section 8
restatement `v2/docs/records/l4e9/L4E9-SECTION8-SET30.draft.md` at `fnd/l4e9s8` f47d1fc4 ("s8" below: blocks 8 and 8a to 8g, its
sections A to D) and the page consistency draft `v2/docs/records/l4e9/L4E9-PAGE-CONSISTENCY-SET30.draft.md` at `fnd/l4e9pc` 8282895e
("PC" below: PC-01 to PC-16 and its contradictions C-1 to C-5). Both drafts were written on 7070f106; the page and the register are
unchanged between 7070f106 and bbba3e53, so their line citations hold; the generator's lines after its PINS table moved by two.

**What this is.** The record of every change of set 31, its source item and its class. It designs nothing, consumes no review and
changes no verdict of a check. The criteria's verdict words are the coordinator's (the set 31 brief), written where s8 left
`[COORDINATOR: criterion N]`. Classes as PC defines them: PRESENTATION OR BINDING (the text says what its cited record already says,
or a count, a pin or a regeneration follows from data in the tree) and CLAIM CHANGE (what the page or the register asserts about the
design changes; every one here narrows a claim or states an open state). No figure a record computes was changed; where a printed
figure differs between records both are printed with their bases. Prototype framing: nothing in the kit is built, bought, powered
or measured.

**How it was run.** The generator on this branch alone refuses at its pins of four cascade outputs (l4e10, l4e11, l4e12 and L4-E7's
P0 output) that 2a pinned at the bytes of the coordinator's commit 2b, not yet committed. For the regeneration and the tests only,
those four outputs were placed in the working tree at exactly the pinned digests (aab5ae6b, 1938c400, 31883eca, 28a5b9fd; read from
the coordinator's uncommitted 2b bytes), and restored to this branch's bytes before every commit; no commit of this branch carries
them. The committed `l4e9_power_path.out` (regen_out: replaced, twice byte-identical, every printed pin current) therefore pins 2b's
digests, as 2a's generator already did. Tests: `python3 -u v2/ecad/tools/tests/run.py test_l4e9. test_public_hygiene.` printed
"tests: 68 passed, 0 failed, 0 skipped" (on the base with the same four outputs: 55 passed, 13 failed).

## A. The changes

| # | Change | Files | Source item | Class |
|---|---|---|---|---|
| 1 | Section 8's head: the DESIGN gate stated apart from the DESK handover gate of part 19, the five states stated once, the citation alias table (lines at 7070f106), the criteria table with the coordinator's verdicts (1 CONDITIONAL, 2 FAIL, 3 PASS, 4 PASS, 5 CONDITIONAL) and their bases as the brief gives them, "closes: NO", set 29's inconsistency, what the P0 round changed | page; generator `GATE` (criteria 1, 2 and 5's constraint and overturn texts) | s8 block 8 | CLAIM CHANGE (criterion 2 CONDITIONAL to FAIL; the verdicts the coordinator's) |
| 2 | 8a: D-10, D-16 and D-17 restated; the P0 round's Layer 8 and 9 findings table; the history note over set 27 to 29's paragraphs | page; `DEFECTS` (D-10, D-16, D-17: state, options, resolution; D-16's constraint) | s8 block 8a; PC-01, PC-02, PC-15 | CLAIM CHANGE |
| 3 | 8b: the cell "Who supplies it" of U-01, U-02 and U-04 (the receiving company since part 19); the set 30 paragraph | page; `CHOICES` supplier fields | s8 block 8b | PRESENTATION OR BINDING (the annex's footing) |
| 4 | 8c: the added paragraph; set 29's paragraph split at the coordinator's sentence | page | s8 block 8c (reconciled, B4) | PRESENTATION OR BINDING |
| 5 | 8d: part 19's footing; OW-4's document cell gains P0-7's two drafts (sha256/16 f3adcf9cebc9655d, 43c524c32e68c085, read on this tree) | page | s8 block 8d | PRESENTATION OR BINDING |
| 6 | 8e: the four checks of the P0 candidate as filed, the method ended, cx46's eighteen items and where each is carried; astra-check-l4close-2 kept as history; the proposed heading; output section 28 gains the checks | generator `cons_check2`, `cons_check2_lines` and their data; page | s8 block 8e (A3) | PRESENTATION OR BINDING (verdicts quoted as filed) |
| 7 | 8f: the ledger's classes after cx46, the withdrawn items, the register's own classes recounted, the D-10, D-16, D-17 and U-01 rows, UDC-2's last cell | generator `cons_class_block`, `D_CLASS`, `D_NEXT`, `U_CLASS`, `cons_comparisons`; page | s8 block 8f (A4); PC-09 | CLAIM CHANGE |
| 8 | 8g: the receiving company's task list; set 29's phase 1 tasks restated (P1-1 narrowed to E-1; P1-2 and P1-3 corrected at the desk by record l8r2); set 29's phase 2 lists rendered from the register | generator `cons_supplier_block`, `cons_p1_tasks`; page | s8 block 8g (B4, B5) | CLAIM CHANGE |
| 9 | FAN_OK withdrawn everywhere: D-17's state, resolution and next action; In short; 1c's C05; 1d's IF-10 cells; R-28's change-list text; R-213 WITHDRAWN; IF-10's check label and the FAN_OK order constraint labelled as a withdrawn row (arithmetic unchanged) | generator; page; register | PC-01 (a) to (f) | CLAIM CHANGE; (f) PRESENTATION OR BINDING |
| 10 | D-16 ADDRESSED IN DRAFTS in In short, the exit row, the decisions, section 12; R-189 restated as S4 and S3 (set 29's acceptance kept for the RSENSE1 arrangement only if restored); R-186 WITHDRAWN and out of `KED_ROWS` | generator; page; register | PC-02 | CLAIM CHANGE |
| 11 | Section 6's 1d counts and its defects paragraph; the exit table's D-17 row; section 12's open defects with D-17 | page; generator `cons_exit_defects` | PC-03 | CLAIM CHANGE |
| 12 | R-206 names U101 LM5069MM-1, the latch-off variant; R-206 to R-208's From name record l8p in the tree | register | PC-04 | PRESENTATION OR BINDING |
| 13 | R-159 restated from E11-29's row word for word (in its Acceptance), its Item summarising it; 5d's E11-29 row, In short and section 6's U-04 row at 40.78 K/W without m, the design target and round 13's method; the generator reads E11-29's row from L4-E11's pinned output (`z3m`, `zw`, `r17t`) | register; generator; page | PC-05 | CLAIM CHANGE |
| 14 | R-246, board P's ideal diode (DD-5), in the register, `CHANGE_ORDER`, `ORDER_CONSTRAINTS` and `CHANGE_SCRIPTS`; `G_L8P` names record l8p's one release | register; generator | PC-06 | CLAIM CHANGE |
| 15 | The counts regenerated (In short, 5b); section 11's counts (235 items); dated paragraphs in section 11 and the register; WITHDRAWN in the register's States legend | page; register | PC-07 | PRESENTATION OR BINDING |
| 16 | R-28: K4's off-list without the fans; its acceptance without FAN_OK | register | PC-08 | CLAIM CHANGE |
| 17 | R-225, R-227, R-232, R-238, R-242, R-244 and R-245 classed KNOWN ENGINEERING DEFECT, ASSIGNED to the ledger's RE-2, RE-4, RE-5 to RE-7 and RE-10 (`RE_ROWS`, `RE_TASK`) | generator; register's Class and Next action (the script's rule) | PC-09 | CLAIM CHANGE |
| 18 | R-236 and R-237 with cx46 item 16's conditions (CO-16) | register | PC-10 | CLAIM CHANGE |
| 19 | In short quotes cx45 and cx46 and keeps astra-check-l4close-2 as history | generator `cons_in_short`; page | PC-11 | CLAIM CHANGE |
| 20 | "l9stk's E-1" (R-159), "l4e7's E-1" (R-240), "decision D-16" (section 12) | register; page | PC-12 | PRESENTATION OR BINDING |
| 21 | R-206 to R-208 in one release with R-222, R-244 and R-246 (record l8p's drafts) | register; generator `G_L8P` | PC-13 | PRESENTATION OR BINDING |
| 22 | IF-01's status on D-10's port-level defect; IF-02 and section 12 with P0-7's figures beside the output's | page | PC-14 (reconciled, B6) | CLAIM CHANGE |
| 23 | D-10 as P0-7 states it (E-1, F1 to F4, the lower-source back-feed) in In short, the exit row, section 6 and section 12; route B2 UNSELECTED and WITHDRAWN AS DRAFTED with no owner item in the data and the `OUT_OF_BASELINE` comment | generator; page | PC-15 | CLAIM CHANGE |
| 24 | R-48 and R-190: FIX, CHECK and APPLY record l8r2's desk drafts (R-221; R-190 with R-228), the receiving company's task only if that check refuses them (`DESK_ROWS`); section 6's list and section 12 | generator; register; page | PC-16 | CLAIM CHANGE |
| 25 | R-227's band 6.3518 to 6.9259 A as `l9t5_f01.out` prints it after cx46 | register | s8 section C, C4 | PRESENTATION OR BINDING |
| 26 | The class rule reads WITHDRAWN first (R-213 is a TEST row, R-186 an EVIDENCE row) | generator `cons_classes` | PC-01 (e), PC-02 (e) | PRESENTATION OR BINDING |
| 27 | `l4e9_power_path.out` regenerated | output | all | PRESENTATION OR BINDING |

**The test expectations changed, each with its evidence basis in a comment** (`v2/ecad/tools/tests/test_l4e9.py`): a WITHDRAWN register
row is admitted when it names its withdrawal (the register's R-210 "WITHDRAWN 5 October 2026: FAN_OK is rejected"; L4E7-P0SOL.md
section 5 for R-186); route B2's draft is exempt from the register and change-list completeness checks through the script's
`OUT_OF_BASELINE` (B2-PRESENCE.md; L4E7-P0SOL.md section 4); D-10 reads OPEN with E-1 and F1 instead of set 29's opening words (L4E7-P0SOL.md
section 4; cx46 item 15); the open defects are D-10 and D-17 and D-16 reads ADDRESSED IN DRAFTS with R-240 (L4E7-P0SOL.md section 5;
cx45's summary; cx46 item 2 for D-17) in five places; D-16 is a PHYSICAL UNCERTAINTY (S3 and S4, SUPPLIER-P1-1-P0SOL.md); D-17's next
action may start ASSIGN (cx46 item 2; the ledger's RE-2). No test was removed; each changed assertion still fails on the old state.

## B. The reconciliations (the narrower claim taken where the drafts overlap)

1. **D-16's state.** s8 8a: "CORRECTED IN DRAFT by P0-7" with S3 and S4 PROVISIONAL; PC-02: "ADDRESSED IN DRAFTS", PROVISIONAL on S3.
   Taken: ADDRESSED IN DRAFTS (the page's own word, never RESOLVED, PC C-1) with both S3 and S4 PROVISIONAL and "not independently
   accepted as closing D-16"; class PHYSICAL UNCERTAINTY (s8 A4).
2. **D-17's state.** s8 8a: "PROVISIONAL, REMAINING ENGINEERING"; PC-01: "OPEN: a correction DRAFTED and PROVISIONAL". Taken: OPEN
   (REMAINING ENGINEERING, RE-2) with its correction PROVISIONAL; it keeps criterion 2 from PASS under the gate's own rule.
3. **The P0 rows' classes in 8f.** s8 8f: "the 25 rows R-220 to R-245, none R-241, are all SETTLED WORK" ([REG:314-338]); PC-09: seven
   of them KNOWN ENGINEERING DEFECT. Taken: PC-09; 8f's counts are recomputed from the register after set 31 (SETTLED WORK 138, PHYSICAL
   UNCERTAINTY 78, KNOWN ENGINEERING DEFECT 13, UNCERTAIN DESIGN CHOICE 6), not s8's base counts (142, 79, 7, 6).
4. **8c and 8g against PC's register restatements.** s8 8c and 8g item 2 name the restatements as owed; PC-05, PC-07, PC-08, PC-09,
   PC-16 and s8's C4 make them. Taken: the texts say they are made in set 31 and that R-48 and R-190 stay OPEN, nothing credited.
5. **8g item 4.** s8: TP-E11-29 NOT EXECUTABLE until L4-E9 restates R-159; PC-05 restates R-159. Taken: still NOT EXECUTABLE until
   its quotation and check are re-taken against the restatement and a supplier agrees the fixture requirement.
6. **IF-02's figures.** PC-14 replaces the output's 2.5485 A and 93.5521 W with P0-7's 2.5378 A and 93.5783 W; this record's output
   computes the former on the drafted RSENSE1 sense (out 4). Taken: both printed, each with its basis (no computed figure changed).
7. **R-159.** PC-05 restates it from E11-29's row word for word; set 29's row also carried the block's transfer rule after the owner's
   L4-QR01 and the superseded 34.42 C/W bar, which E11-29's row does not repeat. Taken: E11-29's row plus those kept obligations.
8. **D-17's What and constraint cells.** s8 replaces the constraint with C-ALLTX rev 3's figures (15.5162 and 16.0718 V); the
   script refuses D-17 without Layer 9's round 2 basis (16.214 V) in its constraint and options, and requires every constraint
   figure printed by its output. Taken: set 29's constraint kept; C-ALLTX rev 3's figures carried in the page's State cell.
9. **D-10's and D-16's options.** s8 replaces set 29's text; the script's citation check, the tests and the history rule hold set
   29's analysis. Taken: s8's text first, then "set 29's options, kept as history". s8's "U5 0.956 V resistive at 3.30 uH" is written
   without the figure: L4-E7's pinned sources do not print 0.956 (the citation check refuses it); L4E7-P0SOL.md section 2 does.
10. **Criterion 2's constraint.** s8's text, prefixed by "two material defects are open: D-10 (E-1) and D-17 (RE-2)" and the
    coordinator's list of open remaining engineering, and followed by set 29's other rows (D-13, D-14, D-15 with its status, D-11,
    R-175), which s8 points to by line only.
11. **Set 29's names kept as history.** D-10's state and In short keep "set 29's B6-ENG-1 as P0-7 restates it" and "round 2's 3.30
    uH loop stays WITHDRAWN as a passing floor" (true on L4E7-P0SOL.md section 4: F3 reads at that loop as a reference).
12. **The five states once.** s8 states them in its head and again under the table; set 31 states them once, in the head, beside the
    DESIGN and DESK gates, as the brief asks.

## C. Not reconciled (both citations; this record settles none)

Citations `[ALIAS:N]` are lines at 7070f106 as in the alias table at the head of the page's section 8; TP29 is
`v2/docs/test-procedures/TP-E11-29.md`.

- **R17's design target:** 0.29 K/W in E11-29's row ([E11:500] at 7070f106) against 0.294 K/W in the annex ([ANX:105]) and
  TP-E11-29's table ([TP29:729]); R-159 prints L4-E11's and names the other (PC C-3).
- **Record l8p's one release:** "five drafts" ([BRK:265]) against the register's R-206, R-207, R-208, R-222, R-244 and R-246; the
  exact membership is record l8p's (PC C-5).
- **The case at the cap:** 15.1307 V in the P0 list ([P0L:18]) against 15.1308 V in the F01 output ([F01:145]); the page uses F01's;
  the P0 list is the coordinator's (s8 C4).
- **One identifier, two items:** E-1 in D-14's row and data (record l9stk's junction limit, kept as s8 keeps D-14) against l4e7's E-1
  (D-10); D-06 the decision against D-06 the defect (s8 C8, C9); PC-12 applied only where it names its places.
- **"Completed independently"** ([P11:89]) against the crediting rule of the common brief; read as ADDRESSED IN DRAFTS, PROVISIONAL (PC C-4).

## D. Left out, and why

- **LH-12** (PC-08): `LAYER5-HANDOVER.md` is not this author's file; PC says its owner record restates it.
- **The re-pins:** records l4e10 and l4e11 pin this page's sha256 and l6r2 the register (the coordinator's at the freeze); L4-E9's
  pins of the three l8p copies at 515f6cf2 (PC-04 assigns their re-take to the coordinator; R-206's From now calls them superseded).
- **45.88 K/W outside PC-05's stated places:** 8a's D-14 row and data, the exit table's D-14 row, U-04's choice row, UDC-1's
  comparison and the 8a history paragraph still state set 29's per-FET bar; s8 keeps D-14 and U-04 unchanged and PC-05 names four
  places; the next set restates them from E11-29's row (40.78 K/W without m).
- **R-176 row 3:** L4E7-P0SOL.md section 5 replaces U5's +-0.240 V line by U5 under 10 mV; neither draft carries it (a finding for the next set).
- **The output's alias citations:** section 8's texts keep s8's `[ALIAS:N]` citations (lines at 7070f106, the alias table at the head of
  section 8); the output prints the same texts without the table.

## E. SESSION decisions (under the owner's standing rule of 26 September 2026)

- **E1. The four cascade outputs placed for the regeneration and tests only.** Reason: 2a's generator refuses this branch's committed
  outputs; the brief says the work does not depend on 2b. Reverse: regenerate after 2b lands; the output then reproduces byte for byte.
- **E2. s8's citations kept**, with an alias table bound to 7070f106, rather than converted to section references (s8's fold-in note
  allows either). Reverse: convert at the next set.
- **E3. s8's proposed 8e heading taken** (s8 A3's reversal). Reverse: restore the old heading.
- **E4. R-48 and R-190 under FIX** (CHECK and APPLY the desk drafts), the class's verb, rather than PC-16's bare "CHECK and APPLY".
- **E5. Set 29's options and names kept as labelled history** in D-10 and D-16 rather than deleted (B9, B11). Reverse: delete them
  with the tests that hold them.

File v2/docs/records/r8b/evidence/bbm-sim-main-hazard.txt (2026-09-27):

requirement: lead >= 1.000 us, hold >= 40.000 us
netlist BOX/out/committed-pcb-b-compute.net: 23 gates, 0 Schmitt buffers, 0 RC nodes; hazard model ON
  1 single vote change (corners)                   runs   162  select moves    162  min lead - us  min hold - us  violations 324
      e.g. select BSEL1 moved at 0.000000000 s with enable BOE1_n LOW (last edge None)
      e.g. select BSEL1 moved at 0.000000000 s with enable BOE1_n LOW (last edge None)
      e.g. select BSEL1 moved at 0.000000000 s with enable BOE1_n LOW (last edge None)
  2 vote returns after r (checker's case)          runs  8478  select moves  33912  min lead 0.000 us  min hold 0.001 us  violations 33912
      e.g. select BSEL1 moved at 0.000000000 s with enable BOE1_n LOW (last edge None)
      e.g. select BSEL1 moved at 0.000000000 s with enable BOE1_n LOW (last edge None)
      e.g. select BSEL1 moved at 0.000000000 s with enable BOE1_n LOW (last edge None)
  3 adversary aimed at the circuit's instants      runs   450  select moves   1800  min lead 0.000 us  min hold 0.000 us  violations 2400
      e.g. select BSEL1 moved at 0.000000000 s with enable BOE1_n LOW (last edge None)
      e.g. select BSEL1 moved at 0.000000000 s with enable BOE1_n LOW (last edge None)
      e.g. select BSEL1 moved at 0.000000000 s with enable BOE1_n LOW (last edge None)
  4 random vote waveforms                          runs  3156  select moves  95620  min lead 0.000 us  min hold 0.000 us  violations 98712
      e.g. select BSEL1 moved at 0.000210747 s with enable BOE1_n LOW (last edge None)
      e.g. select BSEL1 moved at 0.000000007 s with enable BOE1_n LOW (last edge None)
      e.g. select BSEL1 moved at 0.000046611 s with enable BOE1_n LOW (last edge None)
  4 random vote waveforms with power-good toggles  runs  1344  select moves  40980  min lead 0.000 us  min hold 0.000 us  violations 40980
      e.g. select BSEL1 moved at 0.000000389 s with enable BOE1_n LOW (last edge None)
      e.g. select BSEL1 moved at 0.000000396 s with enable BOE1_n LOW (last edge None)
      e.g. select BSEL1 moved at 0.000000017 s with enable BOE1_n LOW (last edge None)
TOTAL runs 13590, select moves 172474, violations 176328

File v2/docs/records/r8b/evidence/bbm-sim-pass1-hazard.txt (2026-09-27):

requirement: lead >= 1.000 us, hold >= 40.000 us
netlist BOX/incoming/pass1.net: 34 gates, 6 Schmitt buffers, 6 RC nodes; hazard model ON
  1 single vote change (corners)                   runs   162  select moves    162  min lead 40.524 us  min hold 0.002 us  violations 162
      e.g. select BSEL1_S moved at 0.000050886 s with the enable off only 50.874 us before and 0.007 us after (required 1.0 and 40.0)
      e.g. select BSEL1_S moved at 0.000086323 s with the enable off only 86.311 us before and 0.006 us after (required 1.0 and 40.0)
      e.g. select BSEL1_S moved at 0.000081578 s with the enable off only 81.569 us before and 0.007 us after (required 1.0 and 40.0)
  2 vote returns after r (checker's case)          runs 14373  select moves  46956  min lead 14.818 us  min hold 0.002 us  violations 47524
      e.g. select BSEL1_S moved at 0.000052486 s with the enable off only 52.474 us before and 0.008 us after (required 1.0 and 40.0)
      e.g. select BSEL1_S moved at 0.000050571 s with the enable off only 50.561 us before and 0.007 us after (required 1.0 and 40.0)
      e.g. select BSEL1_S moved at 0.000048774 s with the enable off only 48.769 us before and 0.004 us after (required 1.0 and 40.0)
  3 adversary aimed at the circuit's instants      runs   450  select moves   1424  min lead 0.005 us  min hold 0.003 us  violations 1464
      e.g. select BSEL1_S moved at 0.000110004 s with the enable off only 109.996 us before and 0.004 us after (required 1.0 and 40.0)
      e.g. select BSEL1_S moved at 0.000110004 s with the enable off only 109.996 us before and 0.004 us after (required 1.0 and 40.0)
      e.g. select BSEL1_S moved at 0.000110004 s with the enable off only 109.996 us before and 0.004 us after (required 1.0 and 40.0)
  4 random vote waveforms                          runs  3110  select moves  15896  min lead 0.007 us  min hold 0.002 us  violations 15910
      e.g. select BSEL1_S moved at 0.000055407 s with the enable off only 2.616 us before and 0.009 us after (required 1.0 and 40.0)
      e.g. select BSEL1_S moved at 0.000070862 s with the enable off only 70.796 us before and 0.003 us after (required 1.0 and 40.0)
      e.g. select BSEL1_S moved at 0.000946394 s with the enable off only 47.039 us before and 0.008 us after (required 1.0 and 40.0)
  4 random vote waveforms with power-good toggles  runs  1390  select moves   7344  min lead 0.268 us  min hold 0.002 us  violations 6120
      e.g. select BSEL1_S moved at 0.000109025 s with the enable off only 108.998 us before and 0.005 us after (required 1.0 and 40.0)
      e.g. select BSEL1_S moved at 0.000117843 s with the enable off only 114.101 us before and 0.003 us after (required 1.0 and 40.0)
      e.g. select BSEL1_S moved at 0.000101293 s with the enable off only 101.280 us before and 0.009 us after (required 1.0 and 40.0)
TOTAL runs 19485, select moves 71782, violations 71180

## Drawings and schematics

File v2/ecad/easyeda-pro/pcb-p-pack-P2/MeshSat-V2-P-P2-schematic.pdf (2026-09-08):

## CELL TAPS, GAUGE BQ4050, SENSE AND SUPPLY FILTERS, THERMISTOR 12345

## FUSE, PROTECTION FETS, GATE NETWORKS, TERMINAL ESD, PACK LEADS 1

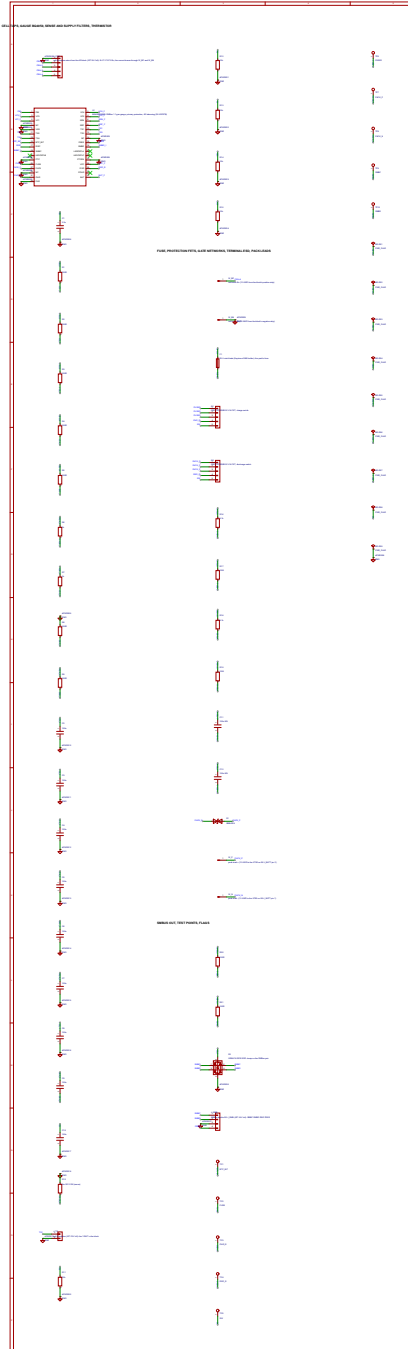
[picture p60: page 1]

J_CELL
cell tap sense wires from the 4S block (JST-XH 1x5): B- C1 C2 C3 B+; the current leaves through W_BP and W_BN

FUSED PACK_P PACK_N SMBC SMBD CELL4 CELL1 CELL2 CELL3 PACK_P PACK_N FUSED SW

BQ4050RSMR: SMBus 1.1 gas gauge, primary protection, 4S balancing (SLUSC67B)

CELL4
cell block B+ (12 AWG from the block's positive strip)

cell block B- (12 AWG from the block's negative strip) ¹ #PWR025

25 A mini blade (Keystone 3568 holder): the pack's fuse

pack lead + (12 AWG to the XT60 on E6 J_BATT pin 2)

pack lead - (12 AWG to the XT60 on E6 J_BATT pin 1)

SMBUS OUT, TEST POINTS, FLAGS

USBLC6-2SC6 ESD clamp on the SMBus pair

J_SMB
SMBus lead to E6 J_SMB (JST-XH 1x4): SMBC SMBD GND PRES

cell thermistor (JST-PH 1x2): the 103AT in the block

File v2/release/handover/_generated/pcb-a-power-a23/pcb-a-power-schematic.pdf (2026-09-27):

J_CP1 | R¹¹⁷ 10k
p15 PACK NODE OVER THE DOCK BLOCK (32.56): | 9 A PINS, PRE-CHARGE, 25 A BLADE, DOCK SIGNAL PINS

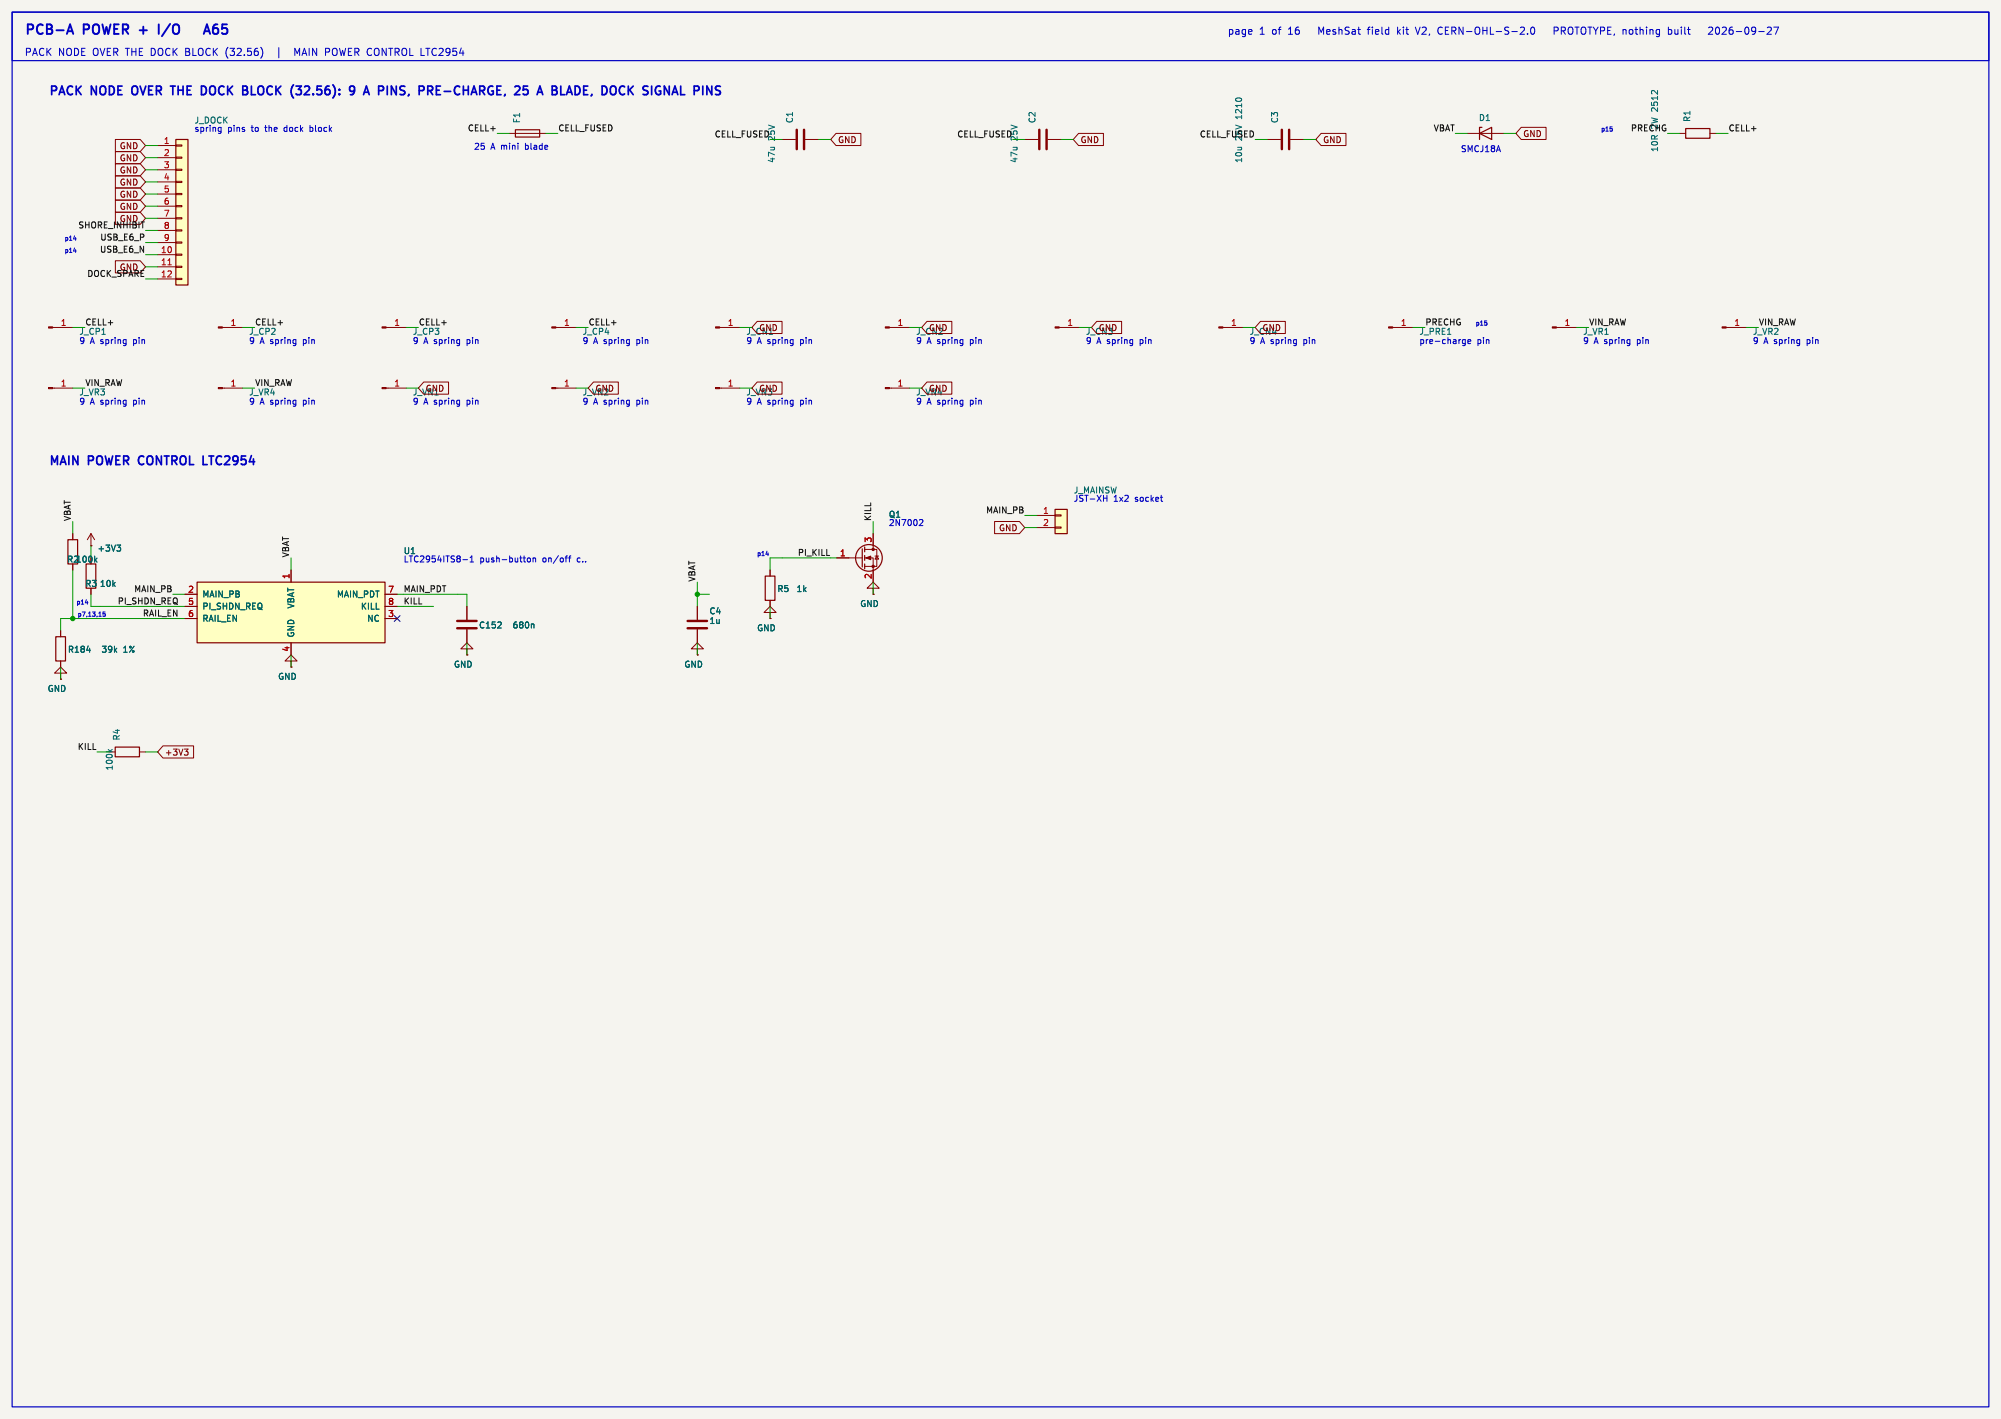
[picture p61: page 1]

GND R¹ 10R ²W ²⁵¹²

J_DOCK
spring pins to the dock block

JST-XH 1x2 socket 9 A spring pin

# J_CP1 R¹¹⁷ 10k

28 U2

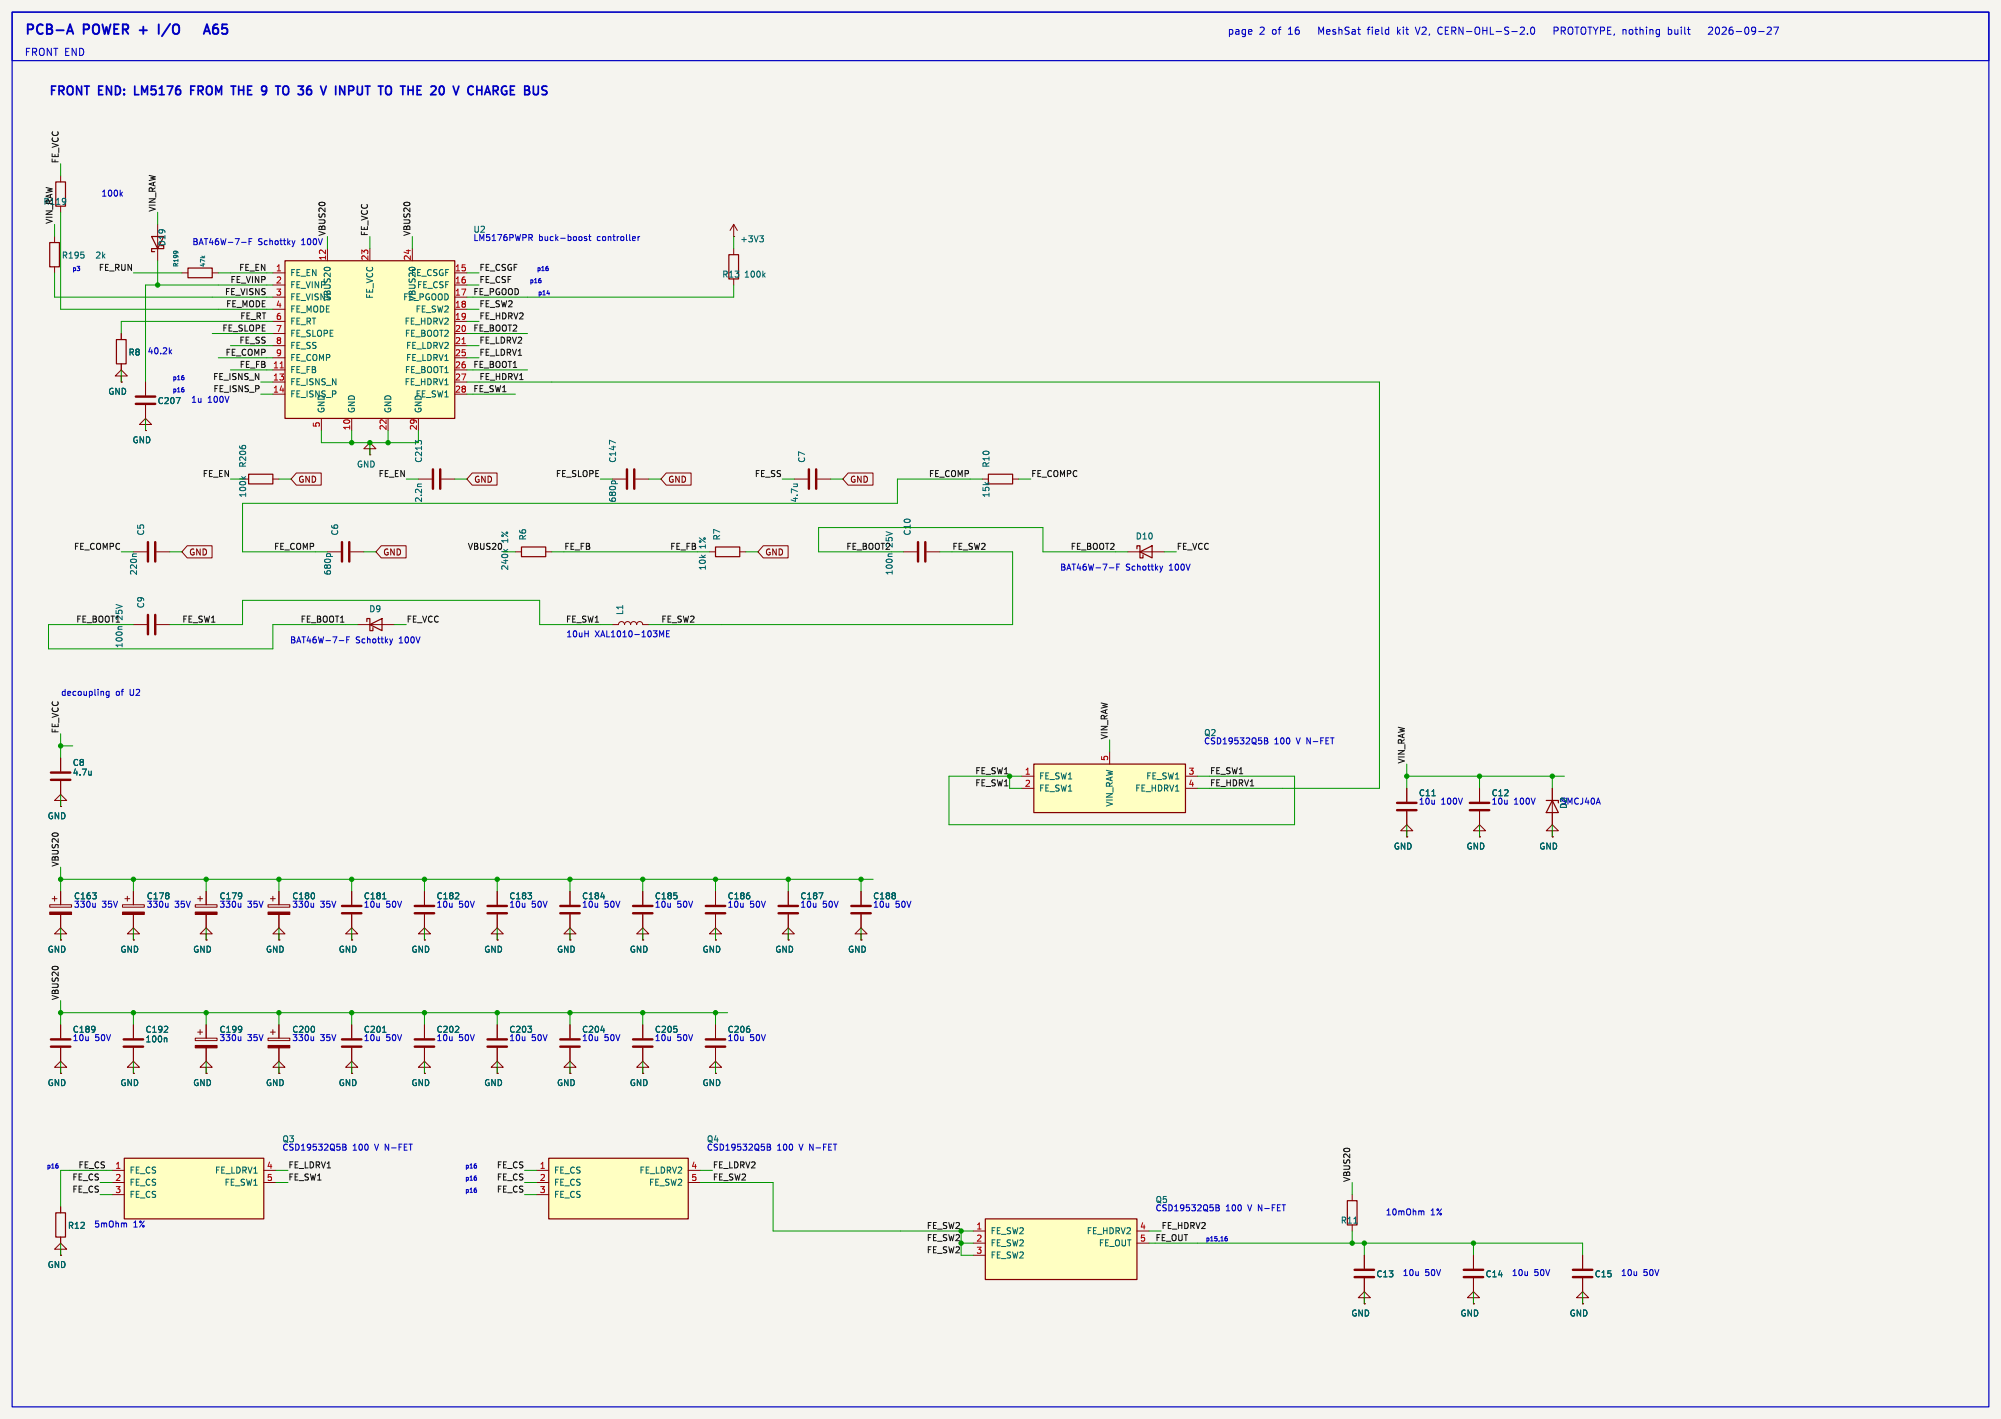
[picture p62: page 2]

FRONT END: LM5176 FROM THE 9 TO 36 V INPUT TO THE 20 V CHARGE BUS

GND R¹ 10R ²W ²⁵¹²

GND | C¹⁷ 100n 25V
R201 | 100k | C¹²⁵ 1n

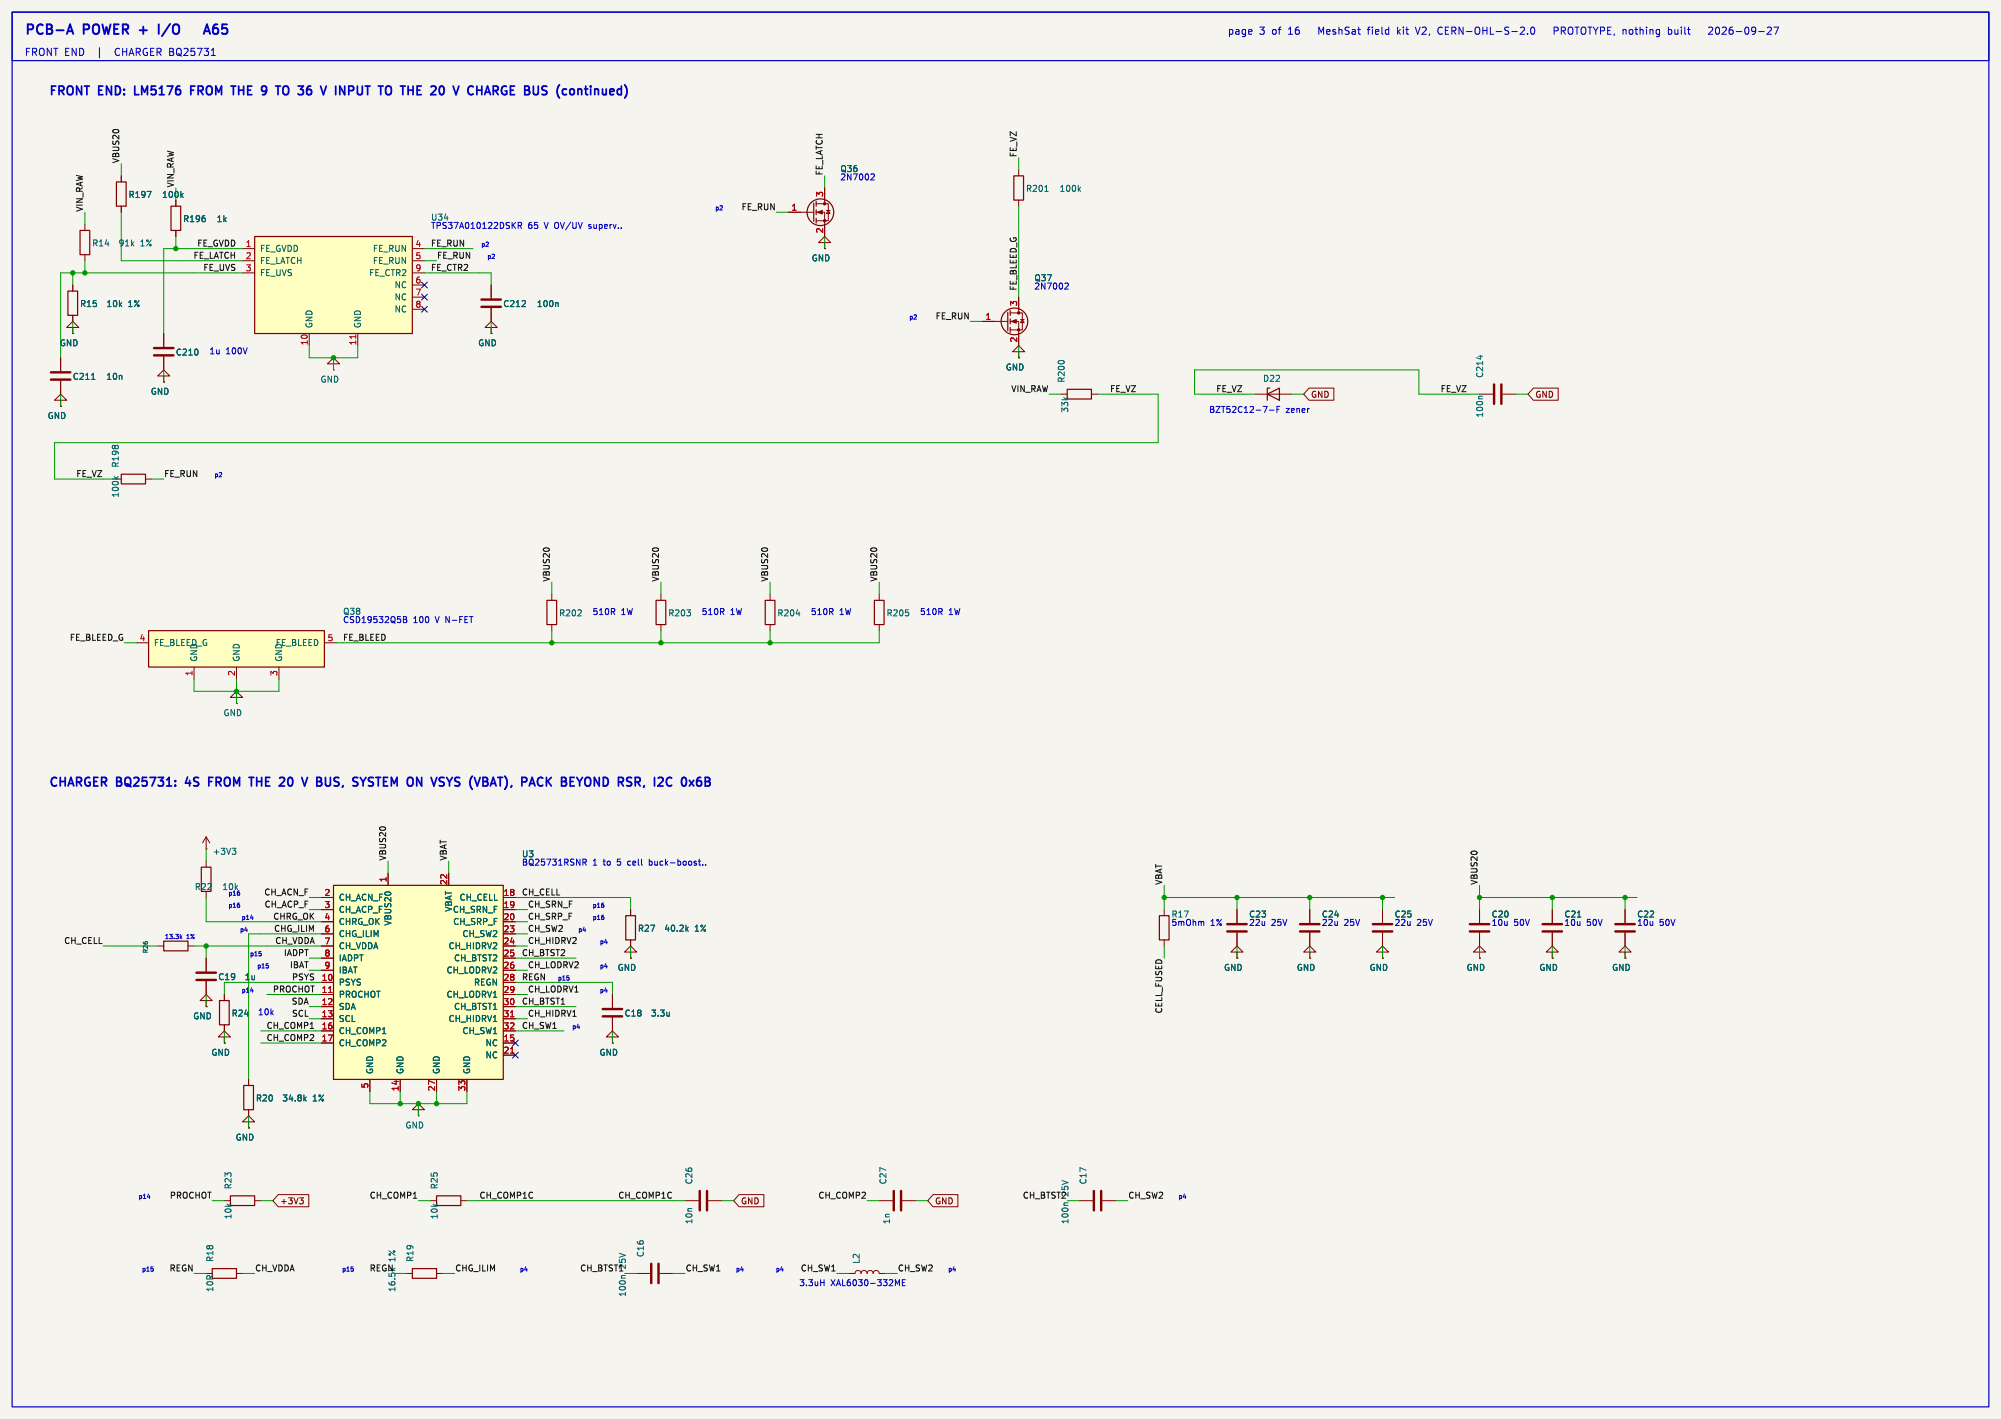
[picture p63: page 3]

GND R¹ 10R ²W ²⁵¹²

GND GND C²¹⁴ 100n R²⁰⁶ 100k

1 GND 14 GND 27 VBAT 22 GND 33 CH_CELL

R201 | 100k | C¹²⁵ 1n

# CH_SW2 CELL+

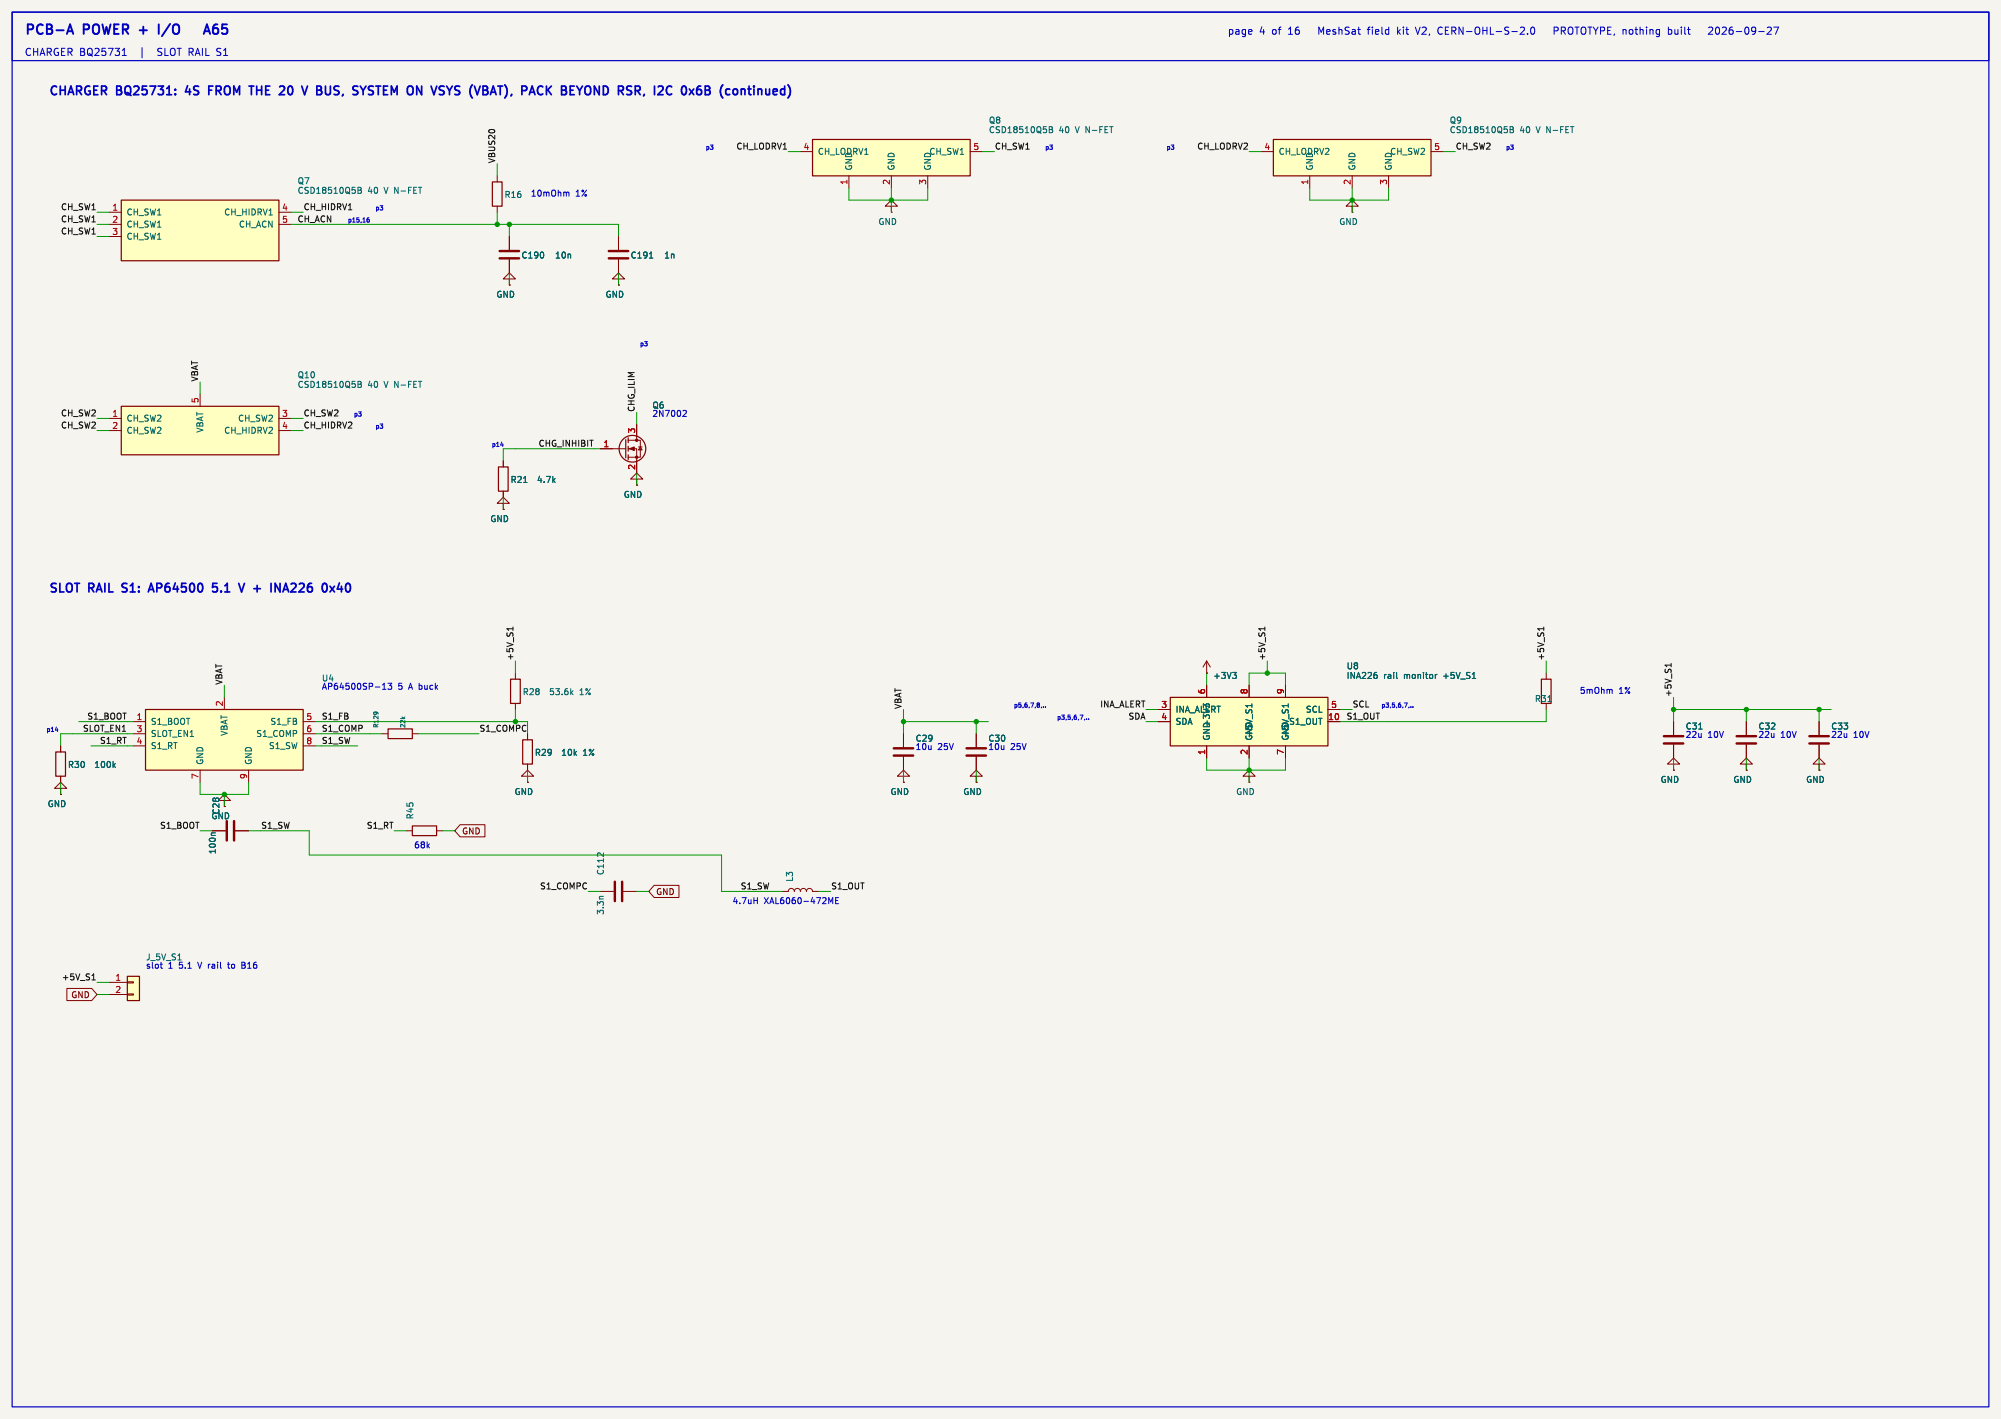
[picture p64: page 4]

GND GND C²¹⁴ 100n R²⁰⁶ 100k

J_CP1 | R¹¹⁷ 10k
R208 | 100k | C⁹ 100n 25V

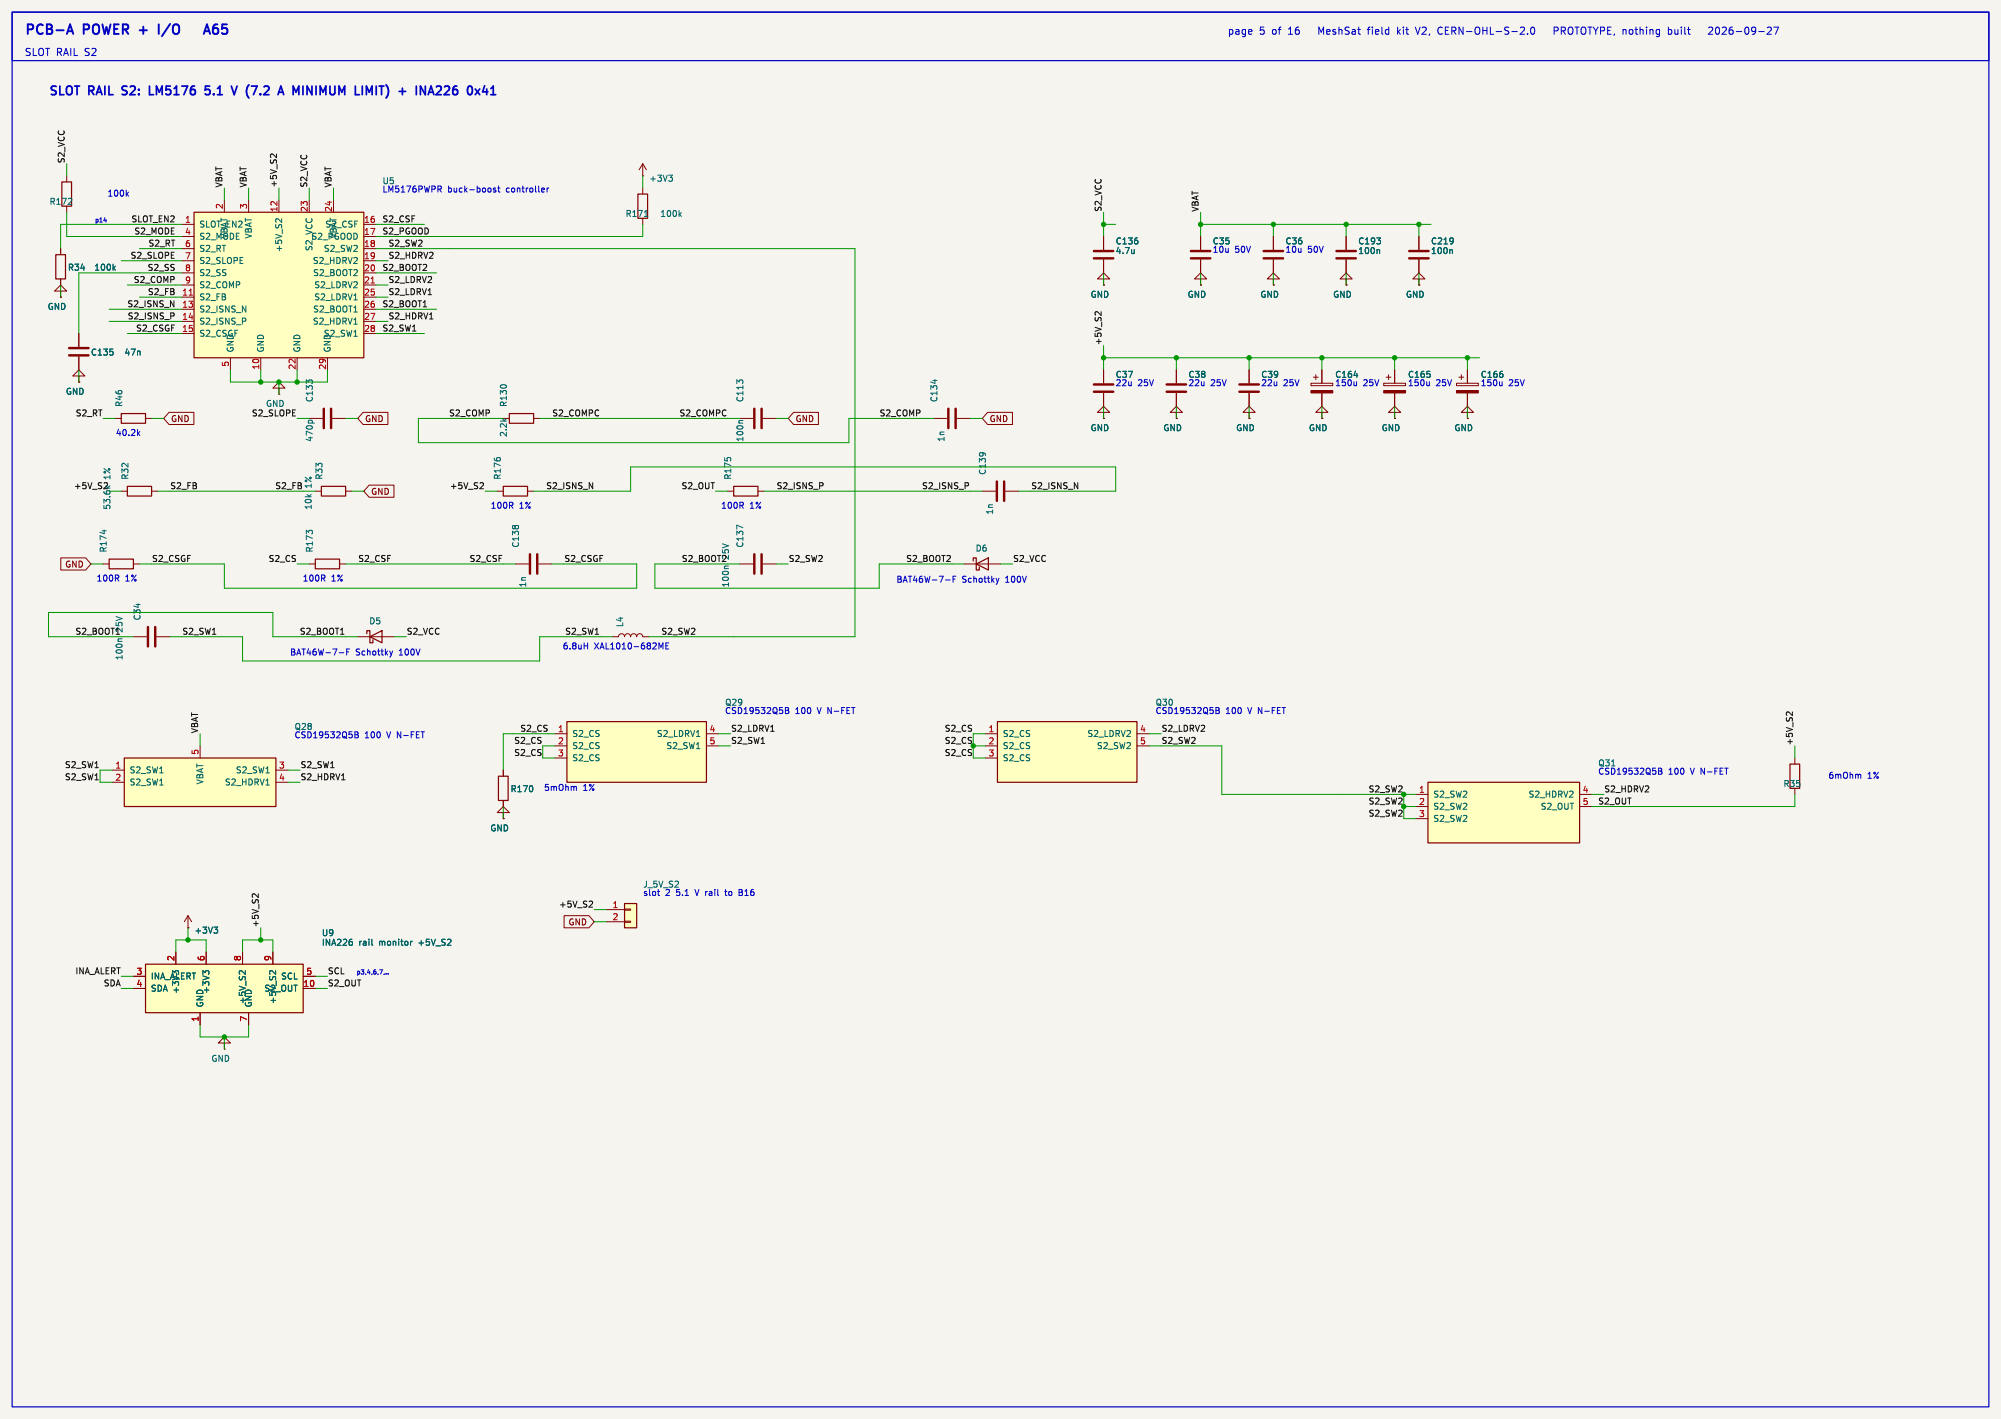
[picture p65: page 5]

GND R¹ 10R ²W ²⁵¹²

p14 SLOT RAIL S2: LM5176 5.1 V (7.2 A MINIMUM LIMIT) + INA226 0x41

3 GND 10 +5V_S2 12 GND 22 S2_VCC 23 GND 29 VBAT 24 S2_CSF 16 S2_PGOOD 17 S2_SW2 18 S2_HDRV2 19 S2_BOOT2 20 S2_LDRV2 21 S2_LDRV1 25 S2_BOOT1 26 S2_HDRV1 27 S2_SW1 28 U5 R80 3.3k

# R37 10k 1% C¹¹⁴ 3.3n

# D10 R¹¹³ 4.7k 1

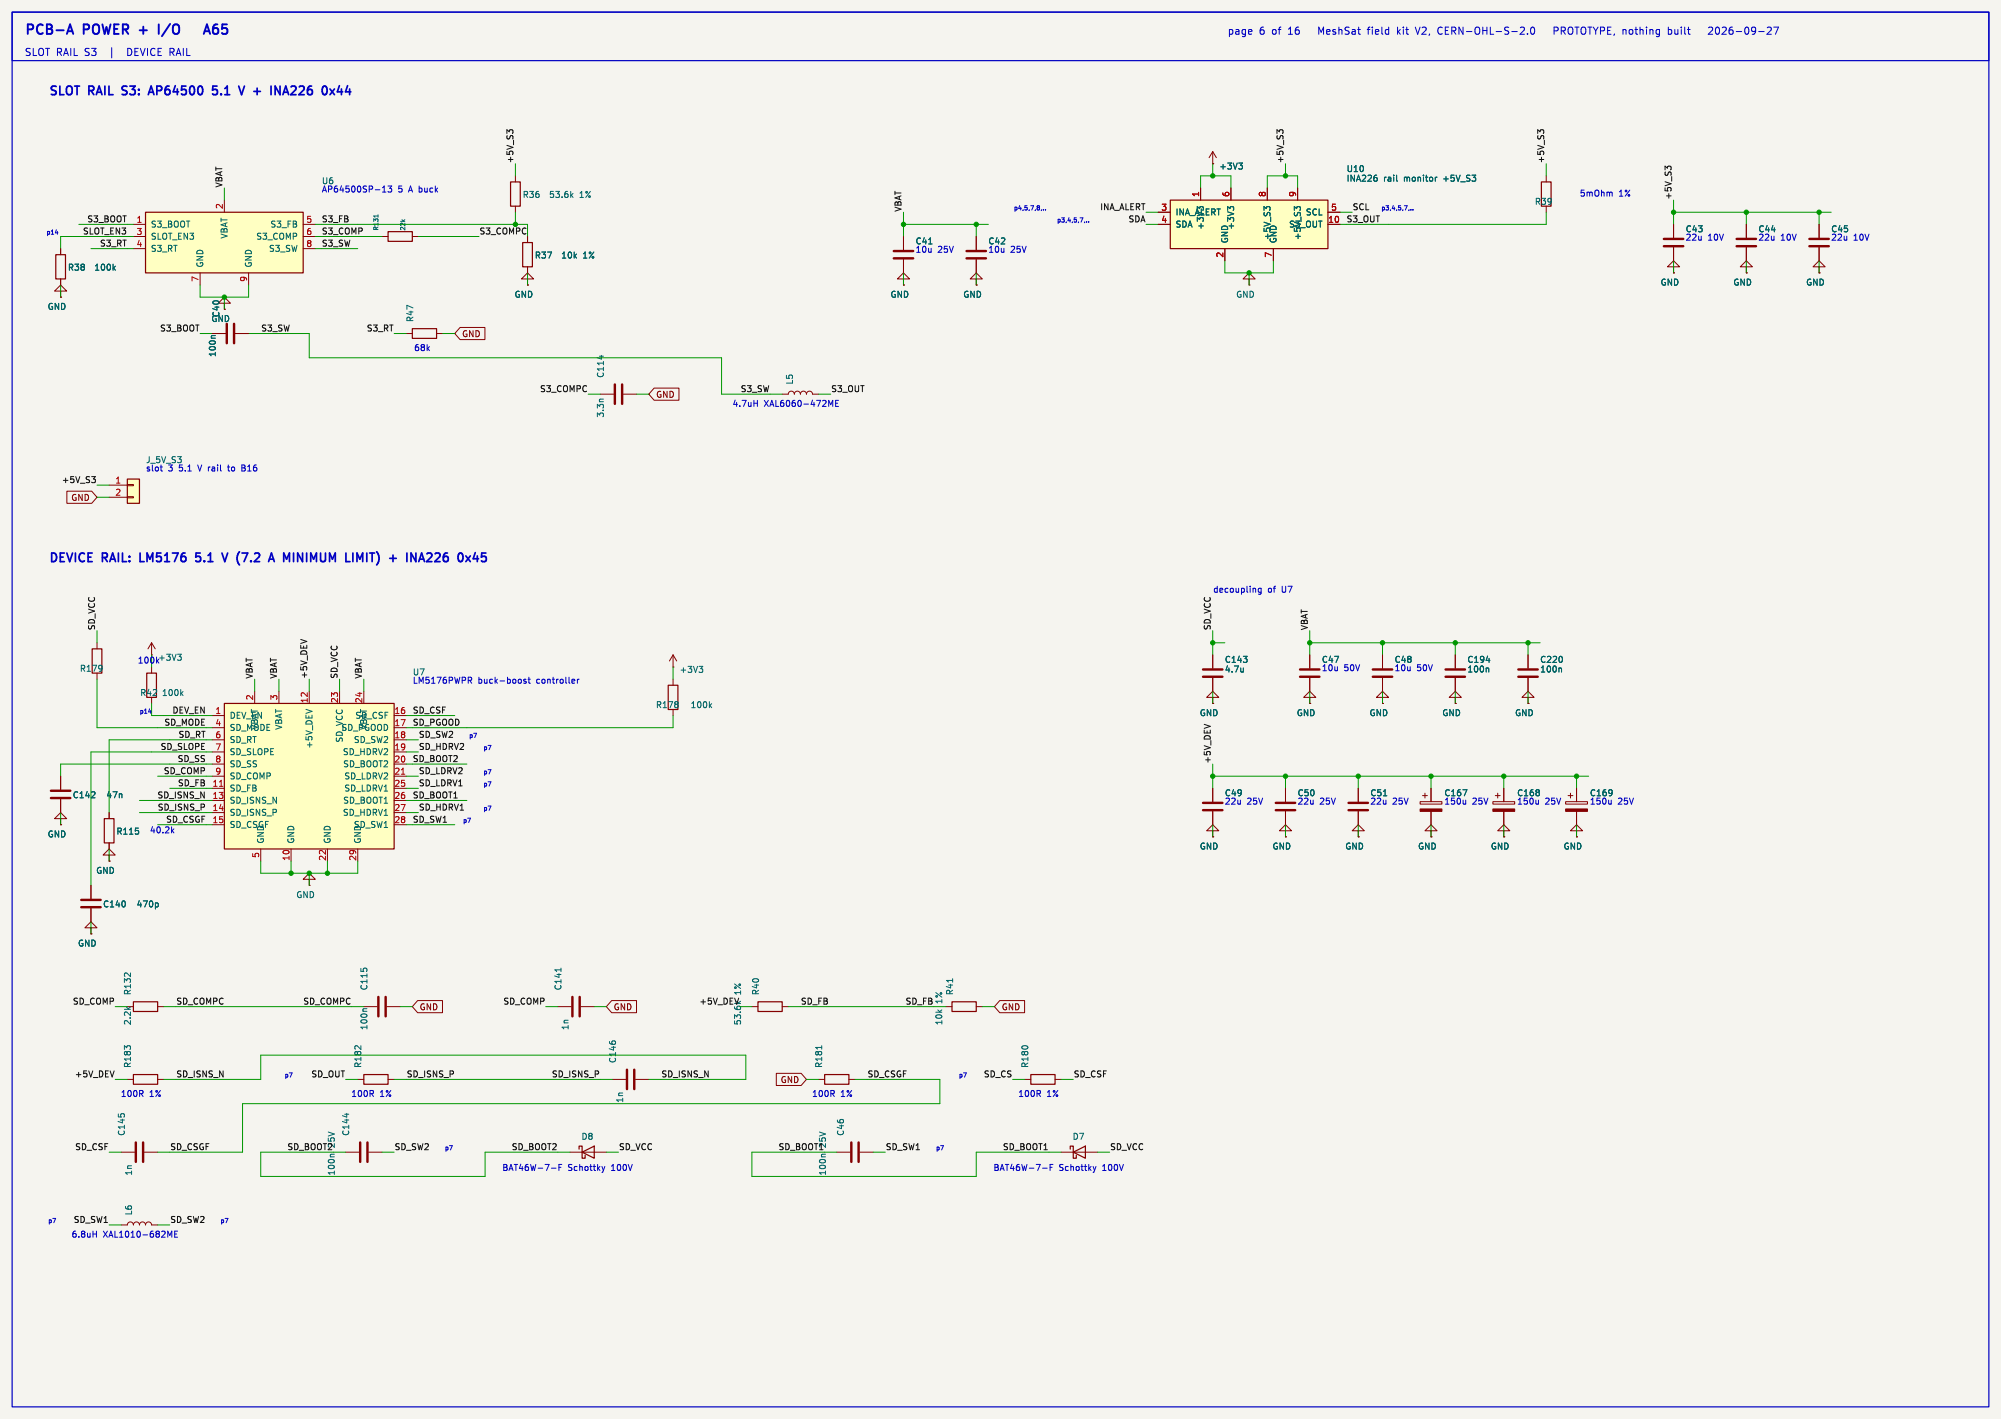
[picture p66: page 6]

GND R¹ 10R ²W ²⁵¹²
USBX_FLT FE_VCC

GND GND C²¹⁴ 100n R²⁰⁶ 100k

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

3 GND 10 +5V_DEV 12 GND 22 SD_VCC 23 GND 29 VBAT 24 SD_CSF

# GND R¹⁸ 10R

# GND R²⁵ 10k GND

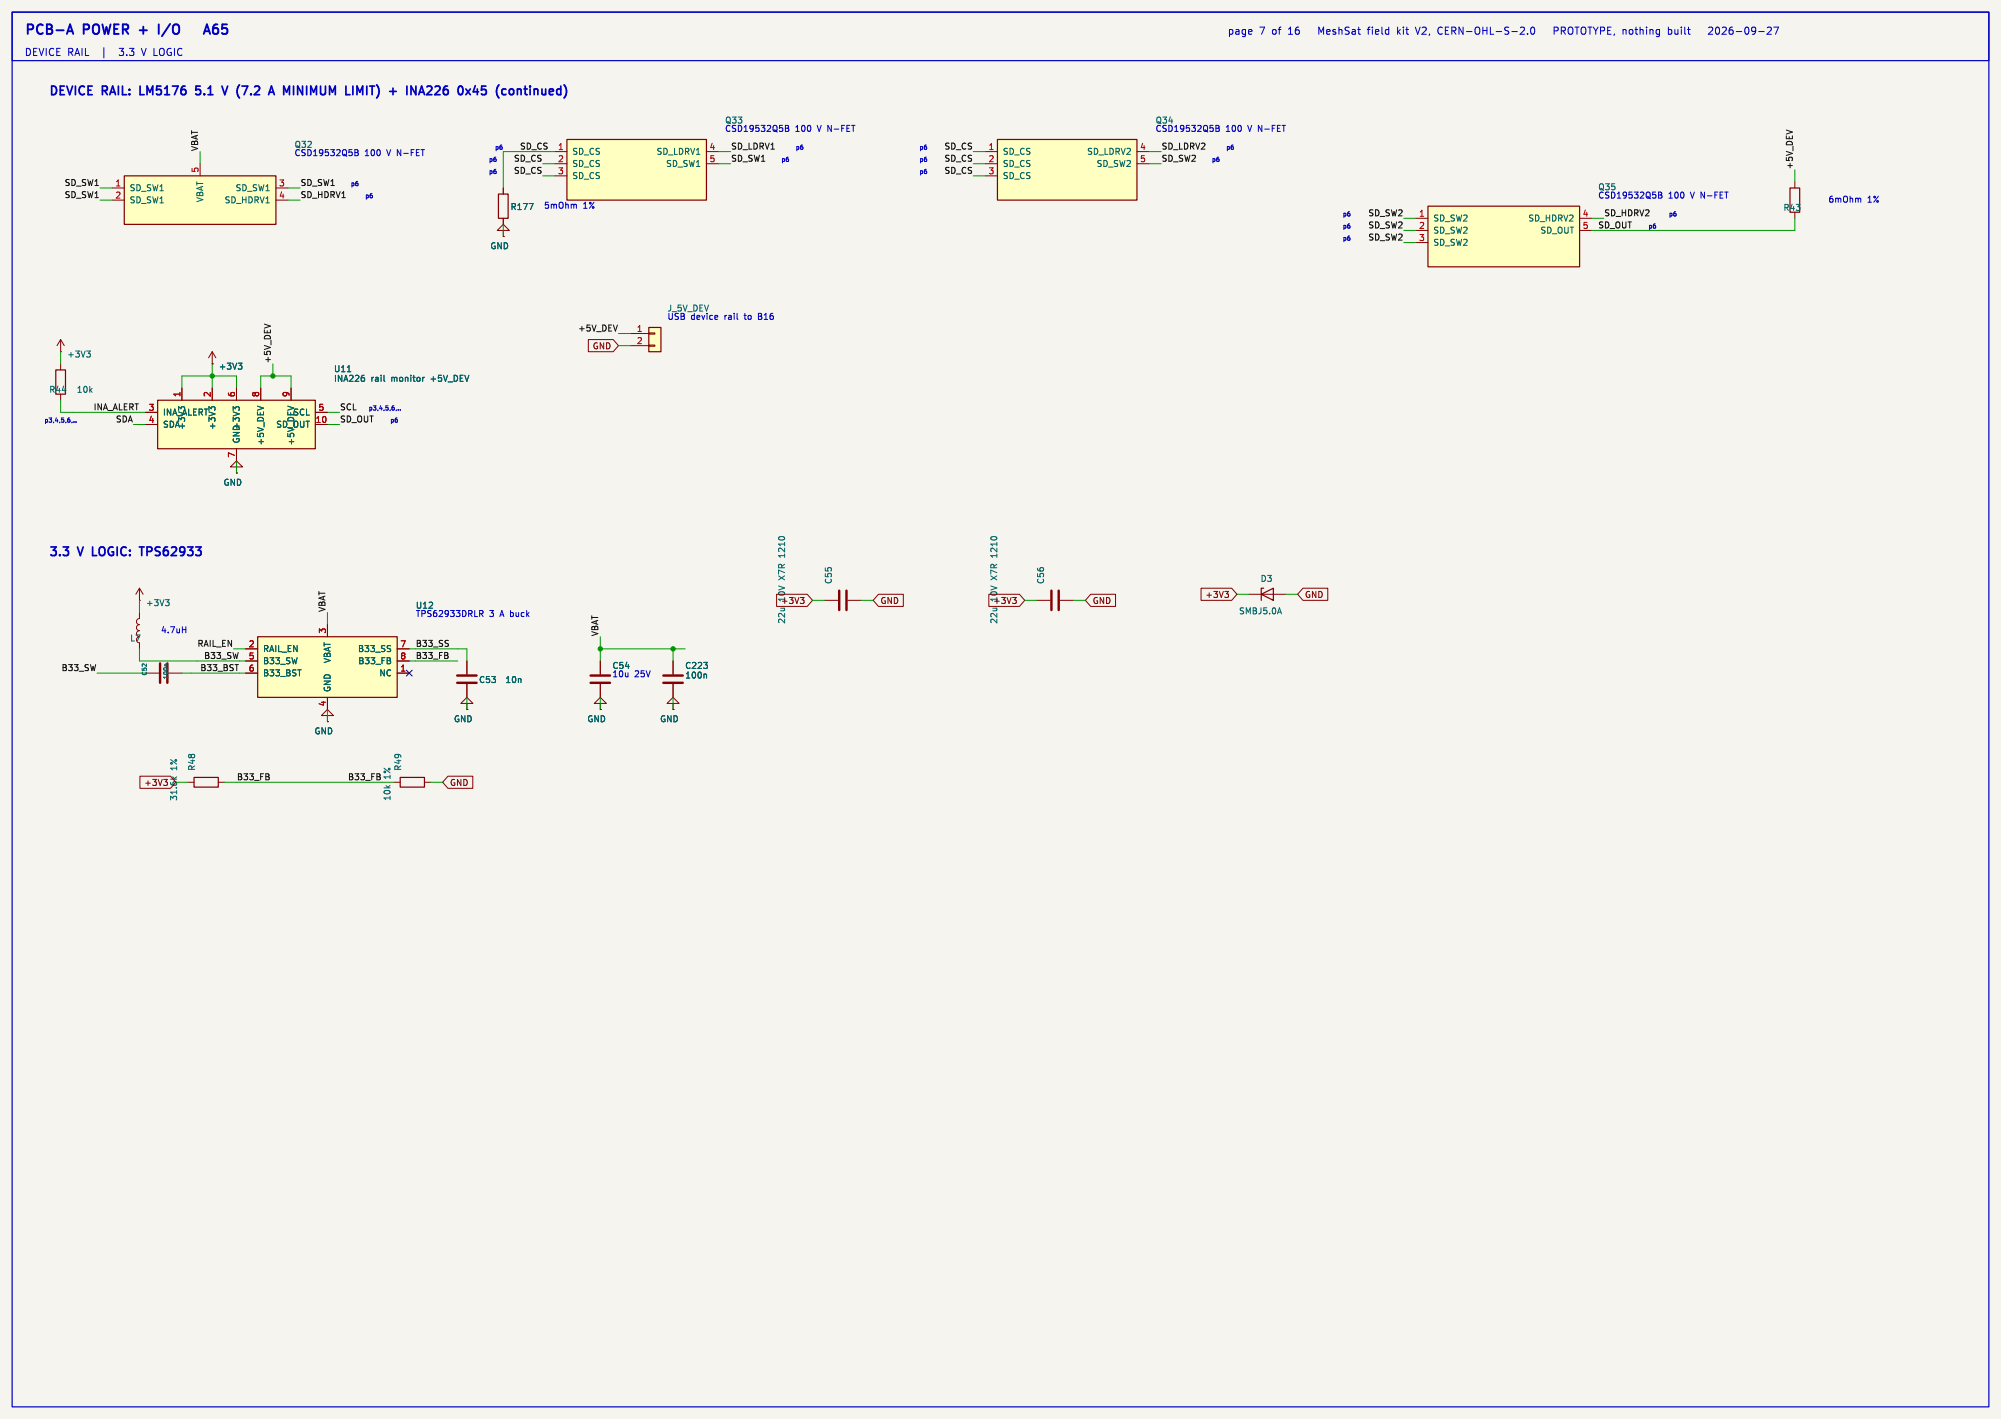
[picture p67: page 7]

GND R¹ 10R ²W ²⁵¹²
CH_SW2 CELL+

GND GND C²¹⁴ 100n R²⁰⁶ 100k

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

J_5V_DEV
USB device rail to B16

R97 GND C⁵⁵ 22u 10V X⁷R ¹²¹⁰

# 15 VBAT

28 U13

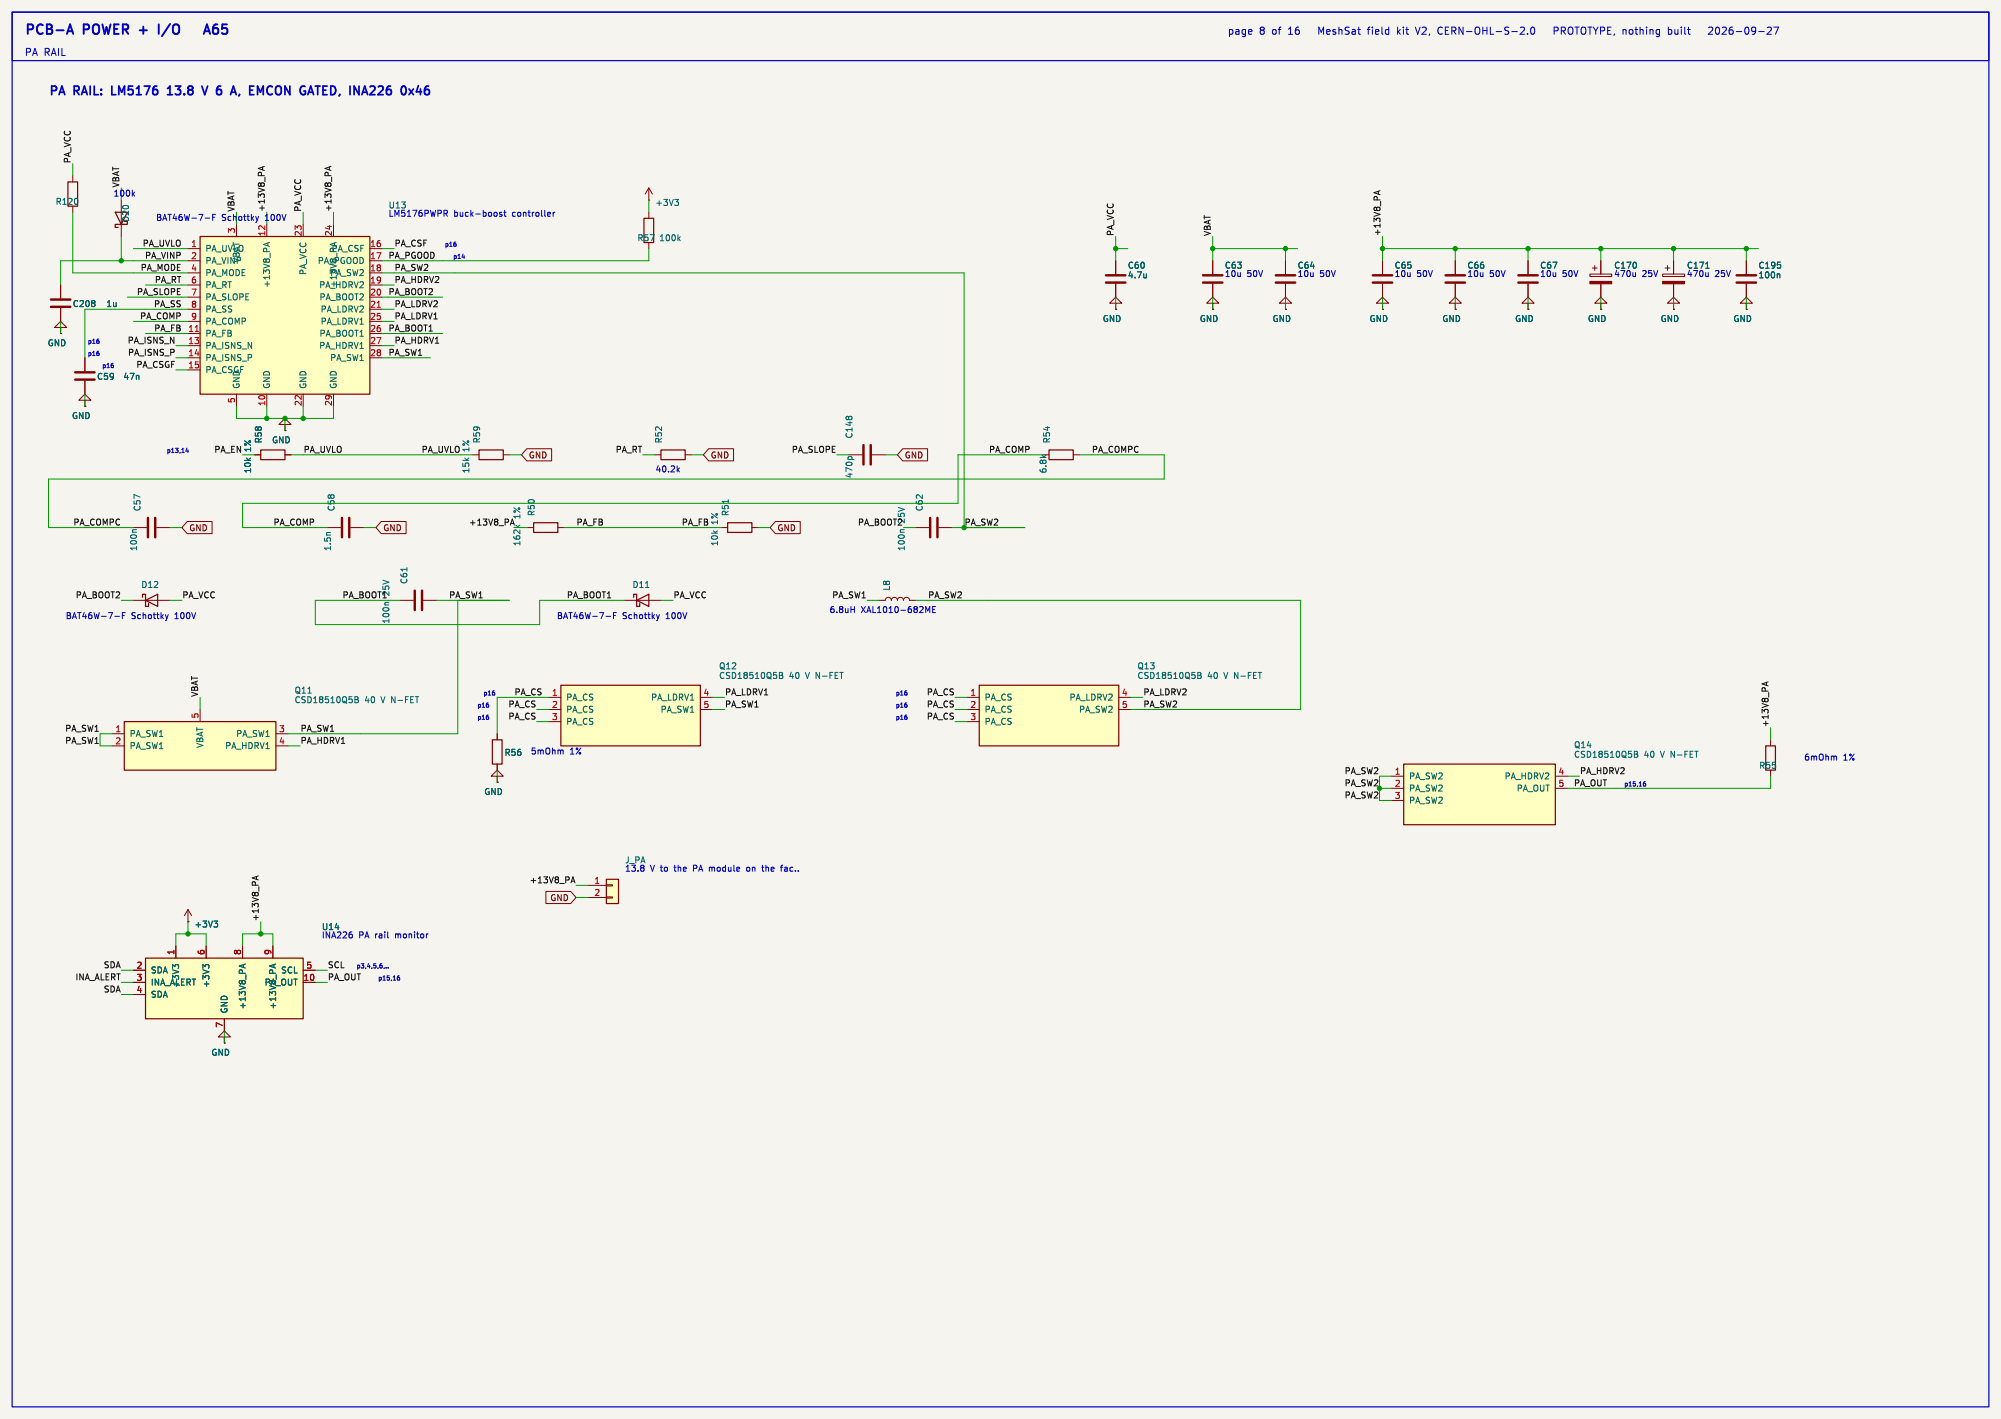
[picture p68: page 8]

GND GND C²¹⁴ 100n R²⁰⁶ 100k

R97 GND C⁵⁵ 22u 10V X⁷R ¹²¹⁰

HF_UVLO 1 HF_VINP 2 HF_MODE 4 HF_RT 6 HF_SLOPE 7 HF_SS 8 HF_COMP 9 HF_FB 11 HF_ISNS_N 13 HF_ISNS_P 14 HF_CSGF 15 VBAT

# GND C¹³³ 470p

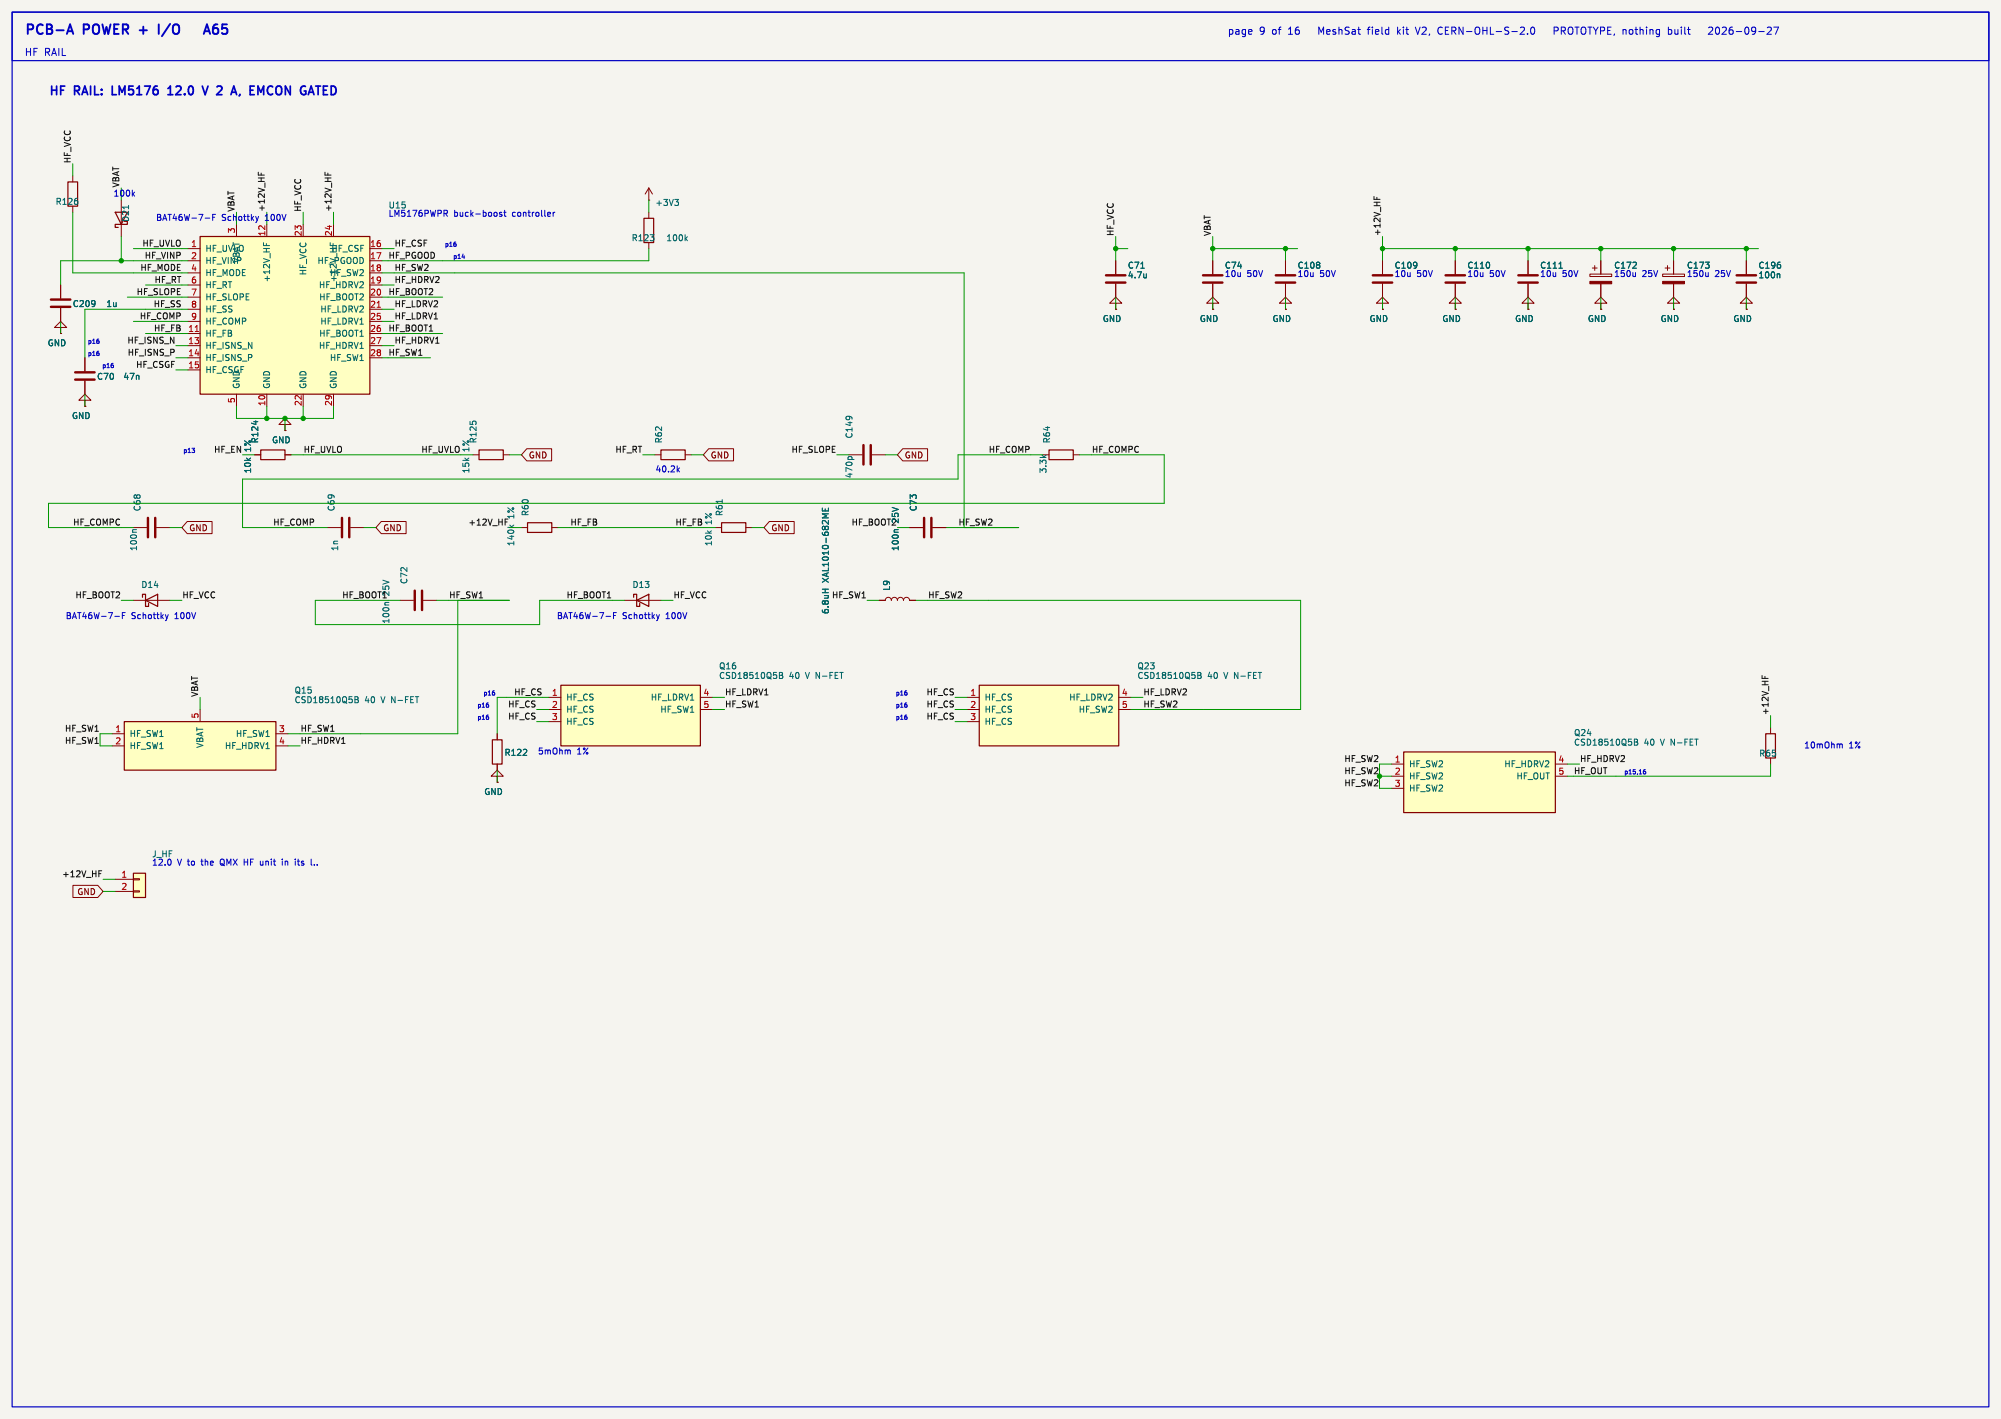
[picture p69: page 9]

GND R¹ 10R ²W ²⁵¹²

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

HF RAIL: LM5176 12.0 V 2 A, EMCON GATED

# D10 R¹¹³ 4.7k 1

R111 | 4.7k | C¹⁰ 100n 25V

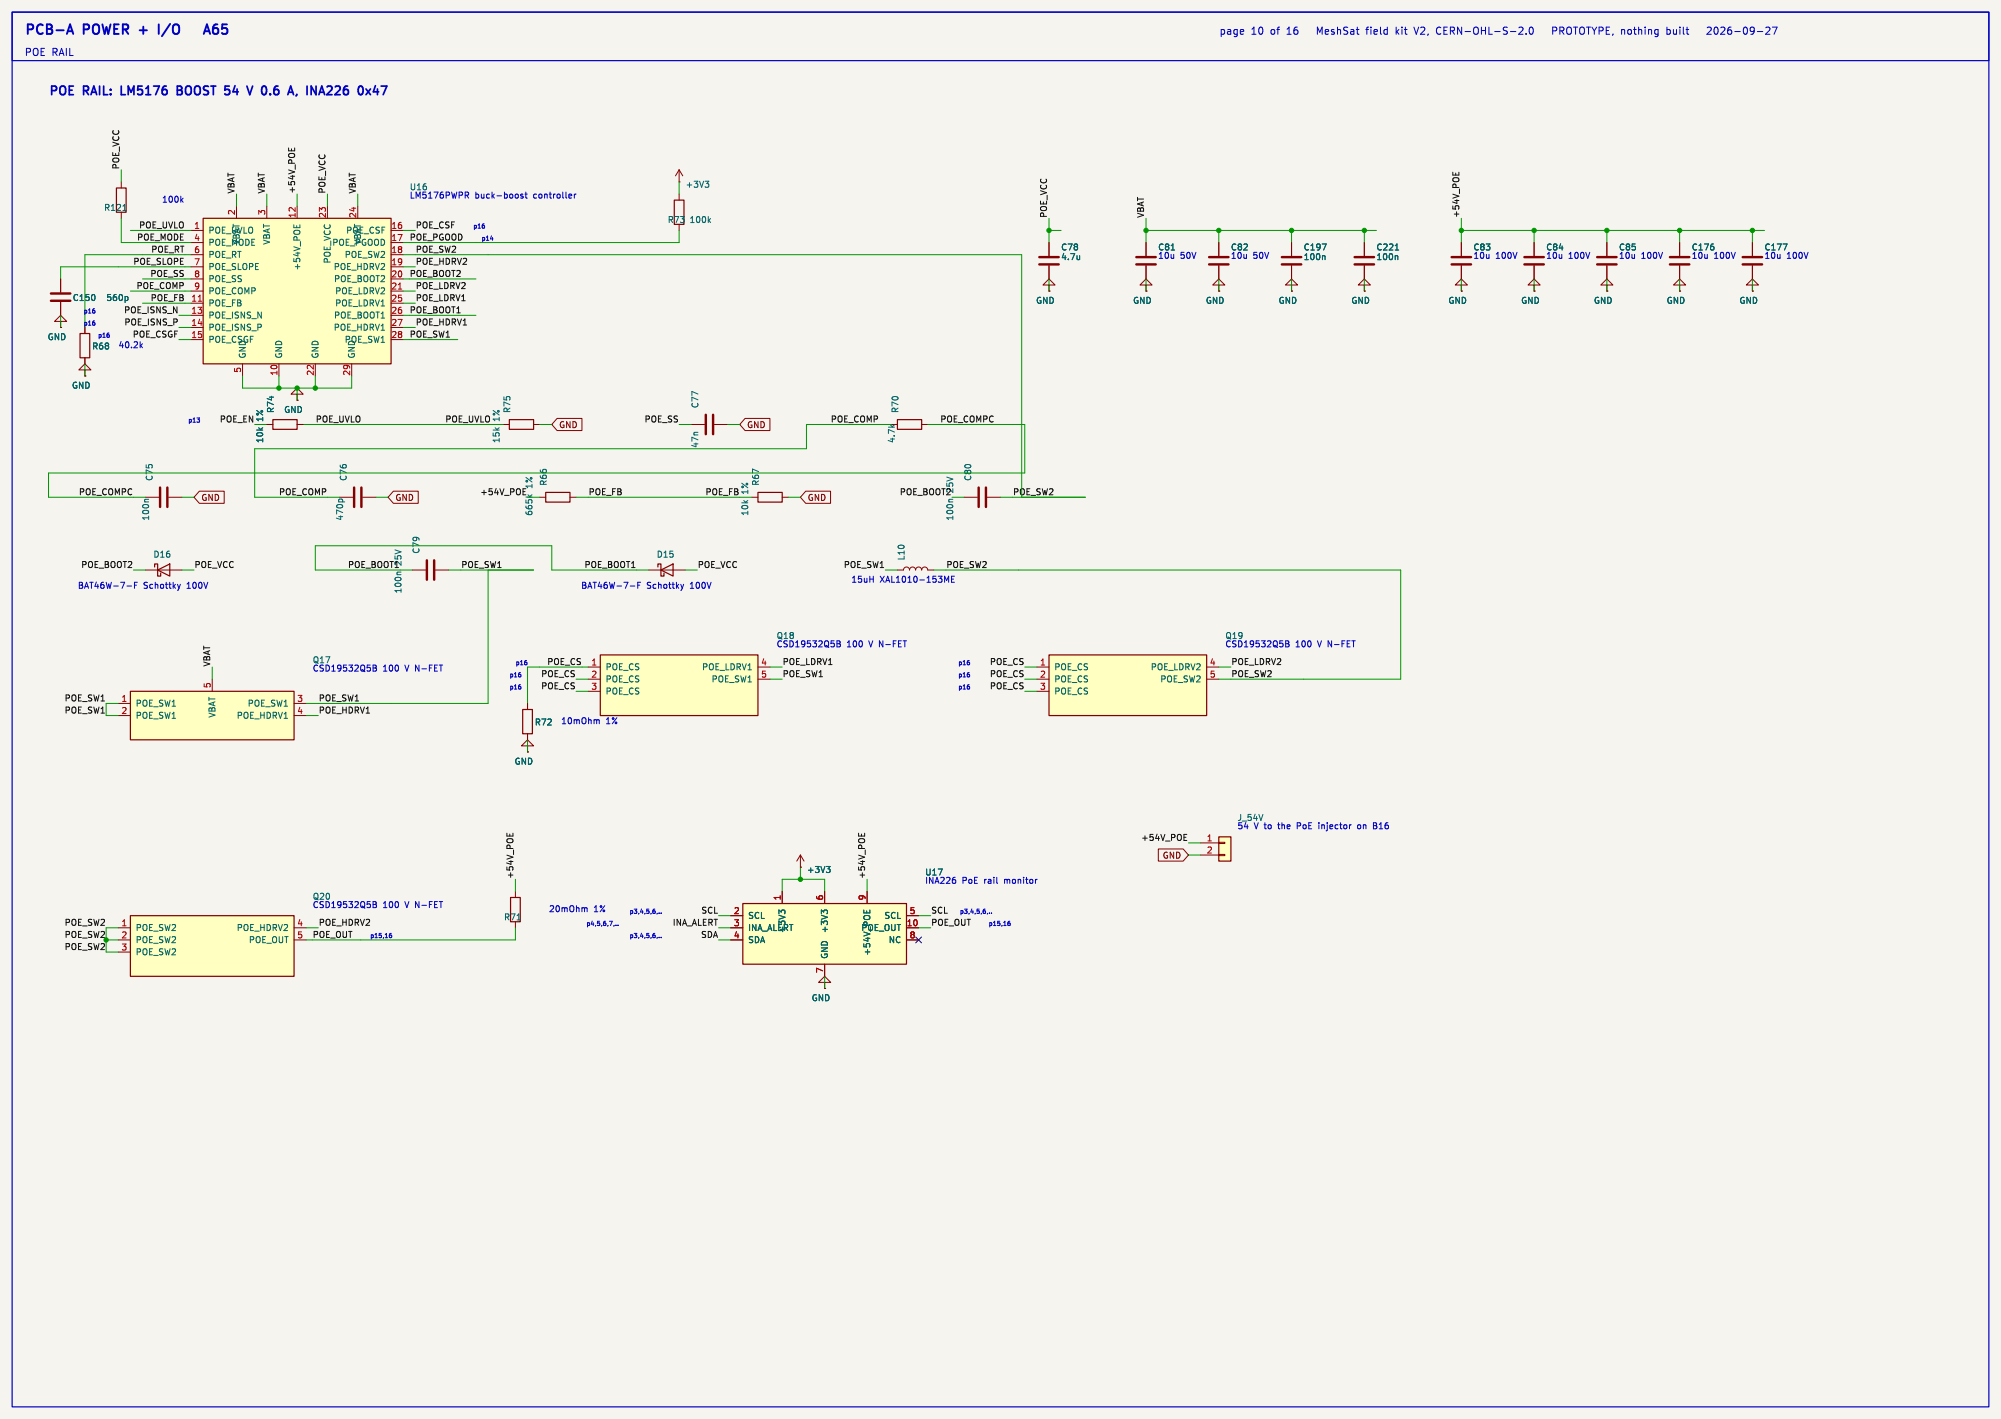
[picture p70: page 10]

GND R¹ 10R ²W ²⁵¹²
USBX_FLT FE_VCC

GND GND C²¹⁴ 100n R²⁰⁶ 100k

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

POE RAIL POE RAIL: LM5176 BOOST 54 V 0.6 A, INA226 0x47

3 GND 10 +54V_POE 12 GND 22 POE_VCC 23 GND 29 VBAT 24 POE_CSF

# GND R¹⁸ 10R

# GND R²⁵ 10k GND

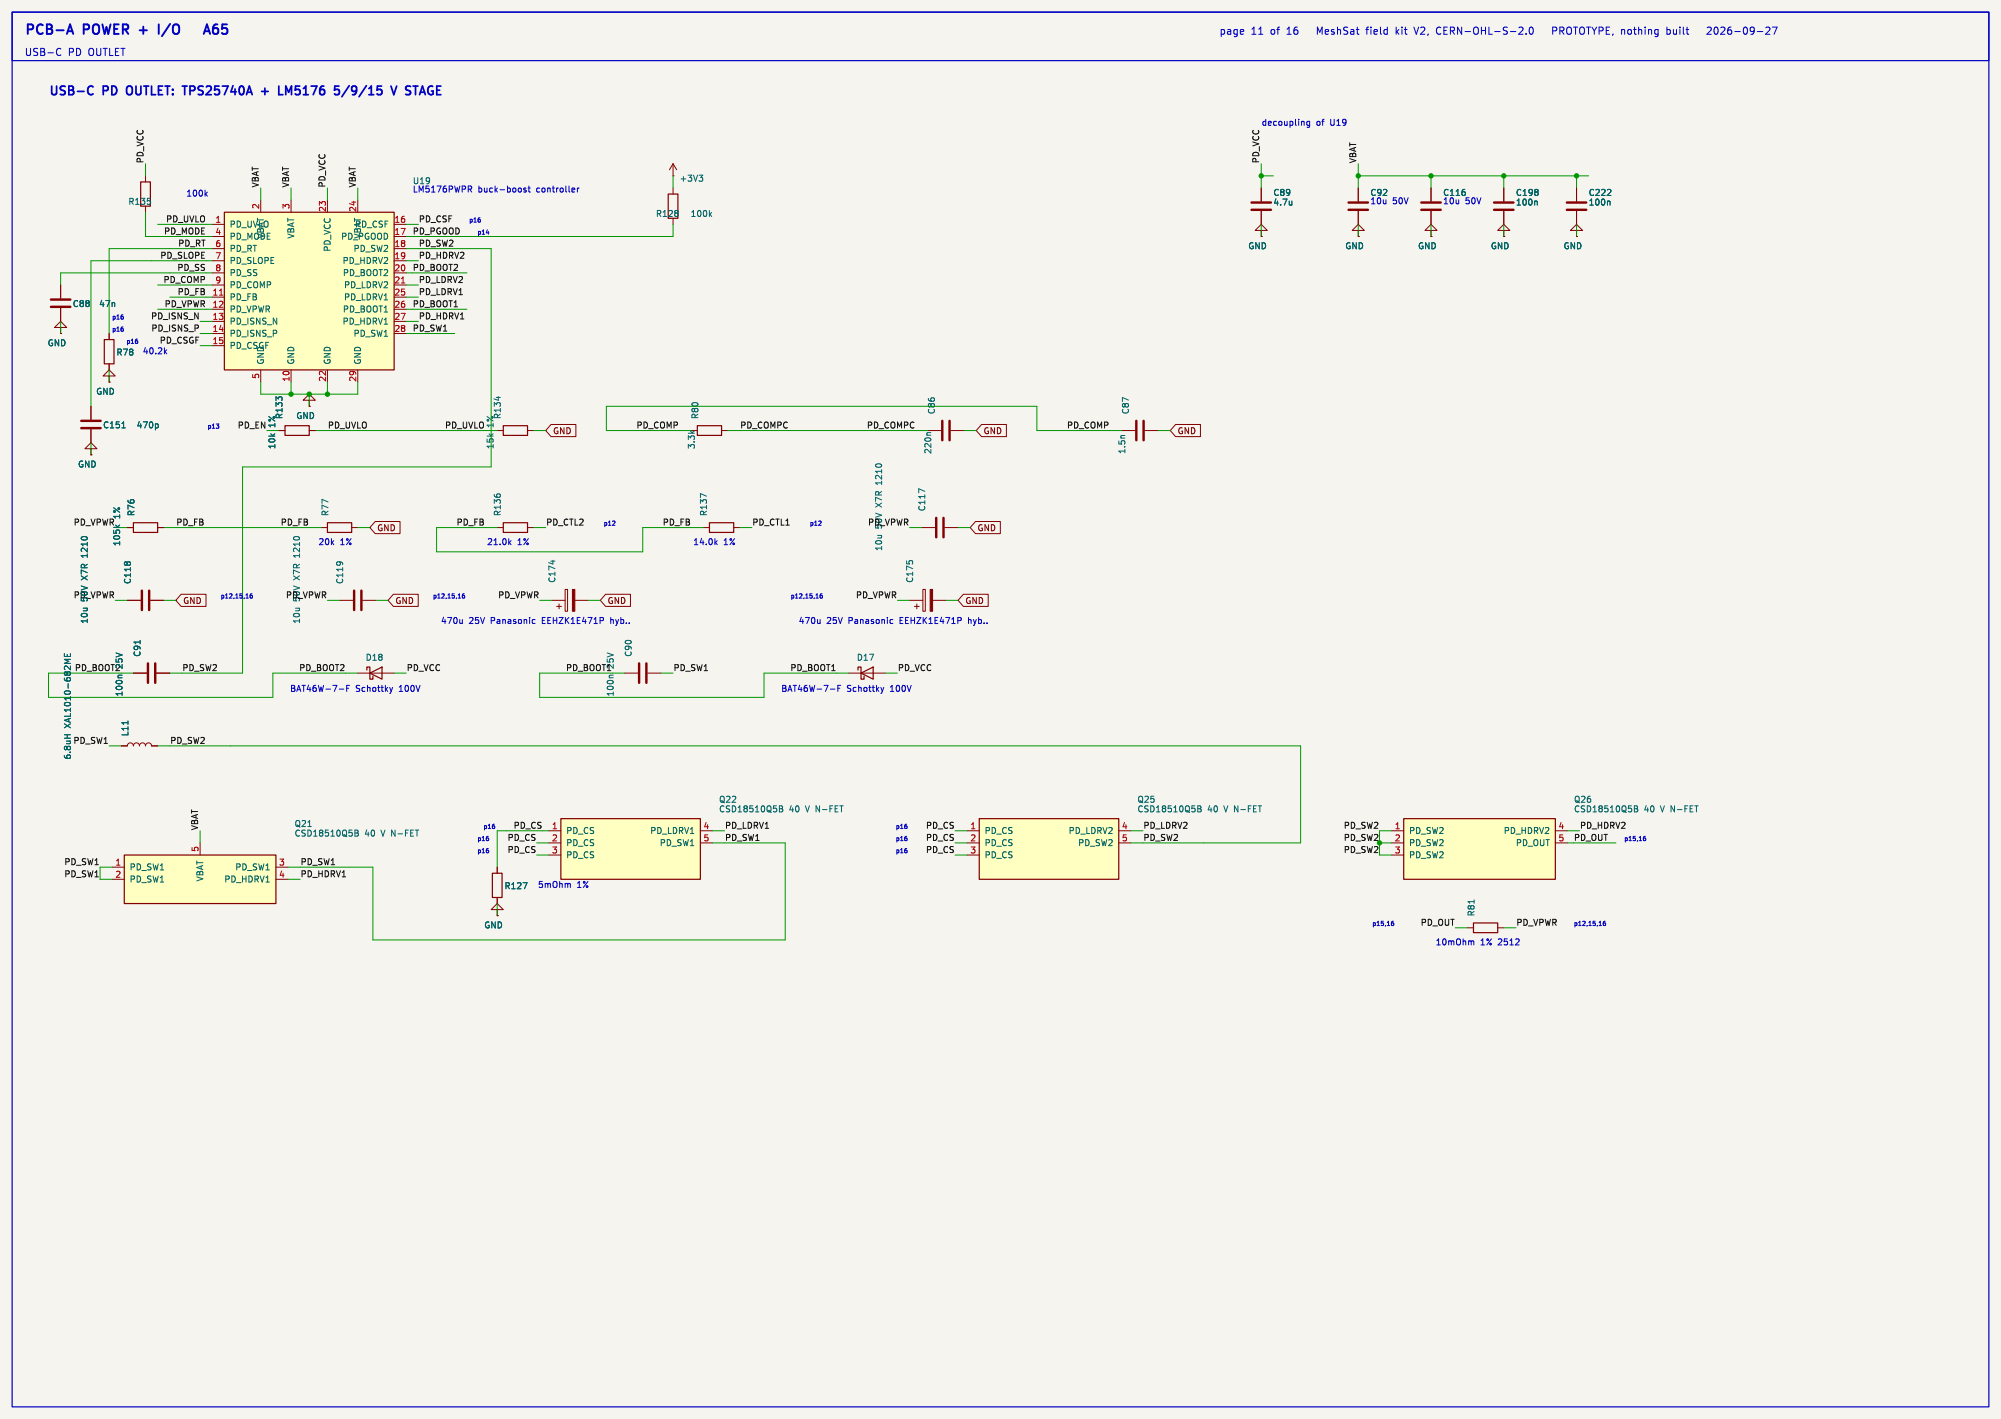
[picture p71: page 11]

GND R¹ 10R ²W ²⁵¹²
CH_SW2 CELL+

GND GND C²¹⁴ 100n R²⁰⁶ 100k

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

R97 GND C⁵⁵ 22u 10V X⁷R ¹²¹⁰

3 GND 10 PD_VCC 23 GND 22 VBAT 24 GND 29 PD_CSF

8 U4 | R¹⁶⁴
R30 100k GND | C¹²⁷ 1n C²⁸ 100n


GND GND C²¹⁴ 100n R²⁰⁶ 100k
PA_COMP PD_VPWR

R97 GND C⁵⁵ 22u 10V X⁷R ¹²¹⁰
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

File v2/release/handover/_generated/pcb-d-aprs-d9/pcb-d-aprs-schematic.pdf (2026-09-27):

# C1 GND R³⁶ 10k

C25 10u | C⁵ 47u 6.3V X⁵R ¹²¹⁰ PA_KEY 2 | +3V³


p7 SA868 EXCITER, UART BRIDGE, T/R RELAY, 10 dB PAD, LPF, PA LEADS, GATE BIAS REGULATOR

# RF_ANT +3V³


2 GND GND GND GND GND

USB HUB TUSB2046I AND ITS 3.44 V LDO, PORT TERMINATIONS, SPARE PORT

GND R¹² | 22
R14 15k R⁴⁹ | 1k


2 GND GND GND GND GND

# C1 GND R³⁶ 10k

# GND GND


USB AUDIO CODEC PCM2912A, HEADPHONE AMPLIFIER, MIC PREAMP, HEADSET LEADS

INR+ 3 OUTR 5 G1 7 CPN 9 CPP 11 EN 13 SGND 15 PAD 17

7 U8

# USB_D8_N VREF


USB AUDIO CODEC PCM2912A, HEADPHONE AMPLIFIER, MIC PREAMP, HEADSET LEADS (continued)

GND GND

PA FLANGE TEMPERATURE: NTC LEAD AND ADC 0x48 ON THE KIT BUS (PWR-F15)

GND R¹² | 22
R14 15k R⁴⁹ | 1k


PTT AND EMCON LOGIC, PTT MIRROR, LEDS, EXPANDER 0x26 WITH LEVEL STAGES, TEST POINTS, FLAGS PTT AND EMCON LOGIC, PTT MIRROR, LEDS, EXPANDER 0x26 WITH LEVEL STAGES, TEST POINTS, FLAGS

C25 10u | C⁵ 47u 6.3V X⁵R ¹²¹⁰ PA_KEY 2 | +3V³
2N7002 | R²⁸ 1.5k


PTT AND EMCON LOGIC, PTT MIRROR, LEDS, EXPANDER 0x26 WITH LEVEL STAGES, TEST POINTS, FLAGS PTT AND EMCON LOGIC, PTT MIRROR, LEDS, EXPANDER 0x26 WITH LEVEL STAGES, TEST POINTS, FLAGS (continued)

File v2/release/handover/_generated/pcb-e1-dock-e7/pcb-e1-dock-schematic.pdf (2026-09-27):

# F3 R²⁵ 10k

# SMBC CELL+ HS_UVLO


J_SMB
SMBus lead to board P

C12 GND C¹⁸ 470n 25V GND R¹⁴ 100k 1% R²¹

GND
BLOCK LANDS (MIRROR OF A22 J_DOCK) AND THE VIN_RAW POWER PADS (EQ-16) green

PANEL TRACKER: J_SOLAR, F2, LT8705A BUCK-BOOST (FBIN 17.6 V, FBOUT 15.1 V, 202 kHz), ORed INTO THE RAW BUS

J_DCF | C²² 100p C15 4.7u 50V
40 | U5 R⁴⁵ | 100R | C¹⁶ 1n


PANEL TRACKER: J_SOLAR, F2, LT8705A BUCK-BOOST (FBIN 17.6 V, FBOUT 15.1 V, 202 kHz), ORed INTO THE RAW BUS (continued)

C12 GND C¹⁸ 470n 25V GND R¹⁴ 100k 1% R²¹

GND
BLOCK LANDS (MIRROR OF A22 J_DOCK) AND THE VIN_RAW POWER PADS (EQ-16) green

solder lands for the 12 signal wir..

# GND GND

# LED1 R⁵⁵ 1M


J_DCF | C²² 100p C15 4.7u 50V
R52 100k R⁵³ | 10k | GND


SENSORS, WATER ELECTRODES, MONITORS, FANS, HEADERS, LID SWITCH, GEIGER SUPPLY

mixer fan 1 under the plate

J_POD
outside sensor pod on the connecto..

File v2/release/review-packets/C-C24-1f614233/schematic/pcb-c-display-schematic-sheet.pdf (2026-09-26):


RIBBON FROM B16, 5 V, 3.3 V LDO, USB AND BUS ESD, FLAGS

PCA9555PW 0x22 EXPANDERS 0x22 / 0x23, MODE INPUTS, EMCON AND ZEROIZE BUFFERS, STRAPS
SCL

p5 RP2040 PANEL CONTROLLER, FLASH, CRYSTAL, BOOTSEL, BUS PULL-UPS

IOVDD 1 GPIO1 3 GPIO3 5 GPIO5 7 GPIO7 9 GPIO8 11 GPIO10 13 GPIO12 15 GPIO14 17 TESTEN 19 XOUT 21 DVDD 23 SWD 25 GPIO16 27 GPIO18 29 GPIO20 31

LED RAIL, INDICATORS, TX LAMP, SWITCHES AND LEADS

LED RAIL, INDICATORS, TX LAMP, SWITCHES AND LEADS (continued)

TEST/ACK 16 mm momentary

J_MAINSW
MAIN button lead to A22 J_MAINSW

E-PAPER ZIF AND THE PDi BOOST, SOUNDER, LIGHT SENSOR, CAMERA MOUNT

4 U_LIGHT
p1,2,5 Vishay VEML7700 ambient light sensor

STANDOFF SCREWS (GND BOND), TEST POINTS, THE REST

STANDOFF SCREWS (GND BOND), TEST POINTS, THE REST STANDOFF SCREWS (GND BOND), TEST POINTS, THE REST (continued)
H6 H1 GND

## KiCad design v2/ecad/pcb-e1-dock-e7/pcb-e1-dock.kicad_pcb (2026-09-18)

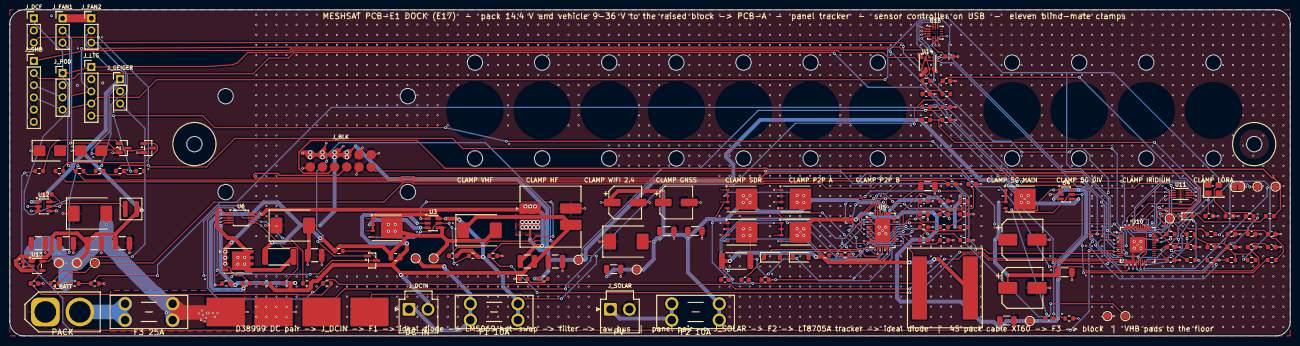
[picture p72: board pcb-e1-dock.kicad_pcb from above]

Board: 4 copper layers, 267.0 x 68.0 mm, 189 parts (0 on the bottom side), 94 nets.

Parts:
C1, C31: 10u 25V 1210; C_1210_3225Metric
C2: 100n 100V; C_0805_2012Metric
C4, C28: 100n 50V; C_0603_1608Metric
C5: 100n (TIMER); C_0603_1608Metric
C6: 1u 100V 1210 (X, input side); C_1210_3225Metric
C7: 1u 100V 1210 (X, bus side); C_1210_3225Metric
C8: 10u 100V X7R 1210; C_1210_3225Metric
C11, C12: 100u 35V Panasonic EEHZK1V101XP hybrid polymer (7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; CP_Elec_6.3x7.7
C13, C14: 10u 50V; C_1206_3216Metric
C15: 4.7u 50V; C_1206_3216Metric
C16: 1n; C_0603_1608Metric
C17, C18: 470n 25V; C_0603_1608Metric
C19: 4.7u 25V; C_1206_3216Metric
C20, C34, C35, C45, C46, C47: 1u; C_0603_1608Metric
C21: 4.7n; C_0603_1608Metric
C22: 100p; C_0603_1608Metric
C23, C30, C38, C39, C40, C41, C42, C43, C44, C48, C49, C50, C51: 100n; C_0603_1608Metric
C24, C25: 39u 35V Panasonic 35SVPF39M polymer (6.9 mm); CP_Elec_8x6.7
C26, C27: 10u 25V; C_1206_3216Metric
C32, C33: 22u 10V X7R 1210; C_1210_3225Metric
C36, C37: 15p; C_0603_1608Metric
D1: SMCJ40A (input surge: 40 V standoff on a line spe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; D_SMC
D2: SMCJ40A (bus clamp: 40 V standoff on the 9 to 36 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; D_SMC
D3: SMCJ18A (pack node clamp); D_SMC
D4: SMCJ28A (panel surge: 28 V standoff, conducting f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; D_SMC
D5: BAT54 boost diode INTVCC -> BOOST1; D_SOD-123
D6: BAT54 boost diode INTVCC -> BOOST2; D_SOD-123
D7: SS14 flyback across fan 1; D_SMB
D8: SS14 flyback across fan 2; D_SMB
F1: 10 A mini blade (Keystone 3568 holder): vehicle i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; Fuseholder_Blade_Mini_Keystone_3568
F2: 10 A mini blade (Keystone 3568 holder): panel inp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; Fuseholder_Blade_Mini_Keystone_3568
F3: 25 A mini blade (Keystone 3568 holder): pack to t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; Fuseholder_Blade_Mini_Keystone_3568
H1, H2: M3 rod pass-through, PCB-A standoff stands here; MountingHole_3.2mm_M3
H3, H4, H5, H6: M3 standoff, raised block; MountingHole_3.2mm_M3
H7, H8: M3, float clamp VHF; MountingHole_3.2mm_M3
H9, H10: M3, float clamp HF; MountingHole_3.2mm_M3
H11, H12: M3, float clamp WIFI 2.4; MountingHole_3.2mm_M3
H13, H14: M3, float clamp GNSS; MountingHole_3.2mm_M3
H15, H16: M3, float clamp SDR; MountingHole_3.2mm_M3
H17, H18: M3, float clamp P2P A; MountingHole_3.2mm_M3
H19, H20: M3, float clamp P2P B; MountingHole_3.2mm_M3
H21, H22: M3, float clamp 5G MAIN; MountingHole_3.2mm_M3
H23, H24: M3, float clamp 5G DIV; MountingHole_3.2mm_M3
H25, H26: M3, float clamp IRIDIUM; MountingHole_3.2mm_M3
H27, H28: M3, float clamp LORA; MountingHole_3.2mm_M3
JP1: BOOTSEL: short while powering to enter the USB bo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; SolderJumper-2_P1.3mm_Open_RoundedPad1.0x1.5mm
J_BATT: Amass XT60-M: the BB-2590/U pack cable BTA-70762-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; AMASS_XT60-M_1x02_P7.20mm_Vertical
J_BLK: solder lands for the 12 signal wires to the block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; PogoTargets_2x6
J_DCF: DCF77 receiver module: 3.3 V, GND, pulse; PinHeader_1x03_P2.54mm_Vertical
J_DCIN: JST-VH socket, 10 A: vehicle and shore DC in 9 to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; JST_VH_B2P-VH_1x02_P3.96mm_Vertical
J_FAN1: mixer fan 1 under the plate (12 V class fan on th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; PinHeader_1x03_P2.54mm_Vertical
J_FAN2: mixer fan 2 under the plate (12 V class fan on th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; PinHeader_1x03_P2.54mm_Vertical
J_GEIGER: Geiger counter module (RadiationD-v1.1 class): 5 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; PinHeader_1x03_P2.54mm_Vertical
J_LTG: AS3935 lightning sensor module (CJMCU-3935 class)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; PinHeader_1x05_P2.54mm_Vertical
J_POD: outside sensor pod on the connector plate (M8 sea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; PinHeader_1x04_P2.54mm_Vertical
J_SMB: pack SMBus (XH or pin header): section A SDA SCL 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; PinHeader_1x06_P2.54mm_Vertical
J_SOLAR: JST-VH socket, 10 A: bare panel in (lead from the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; JST_VH_B2P-VH_1x02_P3.96mm_Vertical
L1: 10uH Coilcraft XAL1510-103MED (Isat 26 A, 10.0 mm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; L_Coilcraft_XAL1510-103
L2: Bourns SRF1260-4R7Y dual-winding choke (7.2 A per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; L_CommonModeChoke_Bourns_SRF1260
L3: 4.7uH XAL4030-472ME; L_Coilcraft_XAL4020-XXX
LED1: green: vehicle input present; LED_0603_1608Metric
LED2: status (GPIO25); LED_0603_1608Metric
PAD_W1: water electrode A (bare copper, +3.3 V through 1 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; SolderPad_8x6
PAD_W2: water electrode B (bare copper, to ADC0); SolderPad_8x6
P_CN: solder pad, 12 AWG wire to the block board return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; SolderPad_8x6
P_CP: solder pad, 12 AWG wire to the block board CELL+ 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; SolderPad_8x6
Q1, Q2: BSC039N06NS 60 V 3.9 mOhm N-FET (PG-TDSON-8: 1-3 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; TDSON-8-1
Q3: BSC028N06NS 60 V 2.8 mOhm N-FET, M1 buck top (TDS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; TDSON-8-1
Q4: BSC039N06NS 60 V N-FET, M2 buck bottom; TDSON-8-1
Q5: BSC028N06NS 60 V N-FET, M3 boost bottom; TDSON-8-1
Q6: BSC039N06NS 60 V N-FET, M4 boost top; TDSON-8-1
Q7: CSD19532Q5B 100 V N-FET (4.6 mOhm at VGS 6 V, Pow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; PowerPAK_SO-8_Single
Q8: 2N7002: SHORE_INHIBIT high pulls UVLO low = input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; SOT-23
Q9: 2N7002 fan 1 low-side switch (1 G, 2 S, 3 D); SOT-23
Q10: 2N7002 fan 2 low-side switch (1 G, 2 S, 3 D); SOT-23
R1, R18, R26: 100k; R_0603_1608Metric
R5: 5 mOhm 1% 3 W 2512 RSENSE (RALEC LR2512-23R005F4); R_2512_6332Metric
R6, R7, R44, R45: 100R; R_0603_1608Metric
R8: 102k 1% (RFBIN1: panel point 17.6 V); R_0603_1608Metric
R9: 7.50k 1% (RFBIN2); R_0603_1608Metric
R10: 115k 1% (RFBOUT1: 15.1 V); R_0603_1608Metric
R11: 10.0k 1% (RFBOUT2); R_0603_1608Metric
R12: 215k 1% (RT: 202 kHz); R_0603_1608Metric
R13, R16, R17, R25, R31, R46, R47, R49, R50: 10k; R_0603_1608Metric
R14, R20, R22, R40, R42: 100k 1%; R_0603_1608Metric
R15: 15.0k 1% (SHDN: enable above about 9.5 V); R_0603_1608Metric
R19: 10mOhm 1% 2512 (hot-swap sense); R_2512_6332Metric
R21: 38.3k 1% (UVLO: 9 V); R_0603_1608Metric
R23: 6.65k 1% (OVLO: 40 V); R_0603_1608Metric
R24: 20k (PWR: power limit); R_0603_1608Metric
R27: 2.2k; R_0603_1608Metric
R28, R33: 1k; R_0603_1608Metric
R29, R30: 27R; R_0603_1608Metric
R32: 1k (BOOTSEL); R_0603_1608Metric
R34, R35, R36, R37: 4.7k; R_0603_1608Metric
R38, R39: 1M; R_0603_1608Metric
R41: 10k 1% (ADC1: 0.091 x bus); R_0603_1608Metric
R43: 22k 1% (ADC2: 0.18 x pack); R_0603_1608Metric
R48: 22R (pulse input series); R_0603_1608Metric
R51: 0R (CSB high: I2C mode; its own net keeps the pin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; R_0603_1608Metric
TP1: DC_IN; TestPoint_Pad_D1.5mm
TP2: DC_P; TestPoint_Pad_D1.5mm
TP3: VIN_RAW; TestPoint_Pad_D1.5mm
TP4: GND; TestPoint_Pad_D1.5mm
TP5: PV_P; TestPoint_Pad_D1.5mm
TP6: TRK_OUT; TestPoint_Pad_D1.5mm
TP7: BLK_SPARE; TestPoint_Pad_D1.5mm
TP8: CELL_F; TestPoint_Pad_D1.5mm
TP9: +5V_E6; TestPoint_Pad_D1.5mm
TP10: SWCLK; TestPoint_Pad_D1.5mm
TP11: SWDIO; TestPoint_Pad_D1.5mm
TP12: E6_RUN; TestPoint_Pad_D1.5mm
TP13: GEIGER_IN; TestPoint_Pad_D1.5mm
U3, U4: LM74700-Q1 ideal-diode controller: 1 VCAP 2 GND 3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; SOT-23-6
U5: LT8705A buck-boost controller, 38-lead QFN 5x7 (p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; WQFN-38-1EP_5x7mm_P0.5mm_EP3.15x5.15mm
U6: LM5069MM-2 hot-swap controller: 9 V on, 40 V off,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; VSSOP-10_3x3mm_P0.5mm
U10: RP2040 sensor controller (USB to B16 through the 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; QFN-56-1EP_7x7mm_P0.4mm_EP3.2x3.2mm
U11: W25Q16JVUXIQ 16 Mbit QSPI flash (USON-8: 1 CS 2 D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; Winbond_USON-8-1EP_3x2mm_P0.5mm_EP0.2x1.6mm
U12: AP63205WU-7 5 V 2 A buck for the controller, the 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; TSOT-23-6
U13: TLV75533PDBVR 3.3 V LDO; SOT-23-5
U14: BME688 inside climate: temperature, humidity, pre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; Bosch_LGA-8_3x3mm_P0.8mm_ClockwisePinNumbering
U15: BMI270 six-axis IMU (I2C 0x68): shock and tilt lo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; Bosch_LGA-14_3x2.5mm_P0.5mm
Y1: 12 MHz ABM8-272-T3 (3225): 1 XIN, 3 XOUT, 2 and 4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; Crystal_SMD_3225-4Pin_3.2x2.5mm

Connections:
/+3V3_E6: C35.1, C38.1, C39.1, C40.1, C41.1, C42.1, C43.1, C44.1, C47.1, C48.1, C49.1, C50.1, J_DCF.1, J_LTG.1, J_POD.1, R25.2, R31.2, R34.2, R35.2, R36.2, R37.2, R38.1, R46.2, R47.2, R49.2, R50.2, R51.1, U10.1, U10.10, U10.22, U10.33, U10.42, U10.43, U10.44, U10.48, U10.49, U11.8, U13.5, U14.2, U14.6, U14.8, U15.5, U15.8
/+5V_E6: C32.1, C33.1, C34.1, J_GEIGER.1, L3.2, TP9.1, U12.1, U13.1, U13.3
/BLK_SPARE: J_BLK.12, TP7.1
/BOOT_J: JP1.1, R32.2
/CELL+: F3.1, J_BATT.2
/CELL_F: C1.1, C31.1, D3.2, D7.1, D8.1, F3.2, J_FAN1.1, J_FAN2.1, P_CP.1, R42.1, TP8.1, U12.2, U12.3
/CELL_MON: R42.2, R43.1, U10.40
/DCF_PULSE: J_DCF.3, R49.1, U10.8
/DCIN_PGD: R25.1, U6.8, U10.15
/DC_F: C4.2, F1.2, Q1.1, Q1.2, Q1.3, R1.2, U3.3, U3.6
/DC_HS: C6.1, L2.1, Q7.1, Q7.2, Q7.3, U6.9
/DC_IN: F1.1, J_DCIN.1, TP1.1
/DC_P: C2.1, D1.2, Q1.5, R19.1, R20.1, R22.1, TP2.1, U3.4, U6.2
/E6_BST: C30.1, U12.6
/E6_DVDD: C45.1, C46.1, U10.23, U10.45, U10.50
/E6_RUN: R31.1, TP12.1, U10.26
/E6_SW: C30.2, L3.1, U12.5
/FAN1_G: Q9.1, R44.2
/FAN1_PWM: R44.1, U10.11
/FAN1_SW: D7.2, J_FAN1.2, Q9.3
/FAN1_TACH: J_FAN1.3, R46.1, U10.13
/FAN2_G: Q10.1, R45.2
/FAN2_PWM: R45.1, U10.12
/FAN2_SW: D8.2, J_FAN2.2, Q10.3
/FAN2_TACH: J_FAN2.3, R47.1, U10.14
/GEIGER_IN: R48.2, TP13.1, U10.9
/GEIGER_PULSE: J_GEIGER.3, R48.1
/GND_V: C2.2, C5.2, C6.2, D1.1, J_DCIN.2, L2.3, Q8.2, R21.2, R23.2, R24.2, U3.2, U6.5
/HS_GATE: Q7.4, U6.10
/HS_OVLO: R22.2, R23.1, U6.4
/HS_PWR: R24.1, U6.7
/HS_S: Q7.5, R19.2, U6.1
/HS_TIMER: C5.1, U6.6
/HS_UVLO: Q8.3, R20.2, R21.1, U6.3
/IMU_CSB: R51.2, U15.12
/IMU_INT1: U10.16, U15.4
/LED_A: LED1.2, R27.2
/LED_STAT: R33.1, U10.37
/LED_STAT_A: LED2.2, R33.2
/LTG_IRQ: J_LTG.5, R50.1, U10.17
/PV_IN: F2.1, J_SOLAR.1
/PV_P: C11.1, C12.1, C13.1, C14.1, C15.1, D4.2, F2.2, Q3.5, R8.1, R14.1, TP5.1, U5.32, U5.33, U5.34
/Q1_G: Q1.4, R1.1, U3.5
/Q2_G: Q2.4, R18.1, U4.5
/QSPI_D0: U10.53, U11.5
/QSPI_D1: U10.55, U11.2
/QSPI_D2: U10.54, U11.3
/QSPI_D3: U10.51, U11.7
/QSPI_SCLK: U10.52, U11.6
/QSPI_SS: R32.1, U10.56, U11.1
/SCL0: J_SMB.2, R35.1, U10.5
/SCL1: J_LTG.4, J_POD.4, J_SMB.4, R37.1, U10.7, U14.4, U15.13
/SDA0: J_SMB.1, R34.1, U10.4
/SDA1: J_LTG.3, J_POD.3, J_SMB.3, R36.1, U10.6, U14.3, U15.14
/SHORE_INHIBIT: J_BLK.8, Q8.1, R26.1, U10.18
/SWCLK: TP10.1, U10.24
/SWDIO: TP11.1, U10.25
/TRK_BG1: Q4.4, U5.14
/TRK_BG2: Q5.4, U5.16
/TRK_BOOST1: C17.1, D5.1, U5.23
/TRK_BOOST2: C18.1, D6.1, U5.17
/TRK_CSN: C16.2, R7.2, U5.2
/TRK_CSP: C16.1, R6.2, U5.3
/TRK_FBIN: R8.2, R9.1, U5.5
/TRK_FBOUT: R10.2, R11.1, U5.6
/TRK_IMONI: R16.1, U5.38
/TRK_IMONO: R17.1, U5.7
/TRK_INTVCC: C19.1, D5.2, D6.2, U5.15, U5.35, U5.36
/TRK_LDO33: C20.1, U5.4
/TRK_LSENSE: L1.2, R5.1, R6.1
/TRK_OUT: C24.1, C25.1, C26.1, C27.1, C28.2, Q2.1, Q2.2, Q2.3, Q6.5, R10.1, R18.2, TP6.1, U4.3, U4.6, U5.29, U5.30, U5.31
/TRK_RT: R12.1, U5.12
/TRK_SHDN: R14.2, R15.1, U5.1
/TRK_SS: C23.1, U5.9
/TRK_SW1: C17.2, L1.1, Q3.1, Q3.2, Q3.3, Q4.5, U5.21
/TRK_SW2: C18.2, Q5.5, Q6.1, Q6.2, Q6.3, R5.2, R7.1, U5.19
/TRK_TG1: Q3.4, U5.22
/TRK_TG2: Q6.4, U5.18
/TRK_VC: C22.1, R13.1, U5.8
/TRK_VCC1: C21.1, R13.2
/U3_VCAP: C4.1, U3.1
/U4_VCAP: C28.1, U4.1
/USB_DM_R: R30.1, U10.46
/USB_DP_R: R29.1, U10.47
/USB_E6_N: J_BLK.10, R30.2
/USB_E6_P: J_BLK.9, R29.2
/VIN_MON: R40.2, R41.1, U10.39
/VIN_RAW: C7.1, C8.1, D2.2, J_BLK.1, J_BLK.2, J_BLK.3, J_BLK.4, L2.2, Q2.5, R27.1, R40.1, TP3.1, U4.4
/WATER_A: PAD_W1.1, R38.2
/WATER_SENSE: C51.1, PAD_W2.1, R39.1, U10.38
/XIN: C36.1, U10.20, Y1.1
/XOUT: C37.1, R28.2, Y1.3
/XOUT_R: R28.1, U10.21
GND: C1.2, C7.2, C8.2, C11.2, C12.2, C13.2, C14.2, C15.2, C19.2, C20.2, C21.2, C22.2, C23.2, C24.2, C25.2, C26.2, C27.2, C31.2, C32.2, C33.2, C34.2, C35.2, C36.2, C37.2, C38.2, C39.2, C40.2, C41.2, C42.2, C43.2, C44.2, C45.2, C46.2, C47.2, C48.2, C49.2, C50.2, C51.2, D2.1, D3.1, D4.1, JP1.2, J_BATT.1, J_BLK.5, J_BLK.6, J_BLK.7, J_BLK.11, J_DCF.2, J_GEIGER.2, J_LTG.2, J_POD.2, J_SMB.5, J_SMB.6, J_SOLAR.2, L2.4, LED1.1, LED2.1, P_CN.1, Q4.1, Q4.2, Q4.3, Q5.1, Q5.2, Q5.3, Q9.2, Q10.2, R9.2, R11.2, R12.2, R15.2, R16.2, R17.2, R26.2, R39.2, R41.2, R43.2, TP4.1, U4.2, U5.11, U5.13, U5.37, U5.39, U10.19, U10.57, U11.4, U11.9, U12.4, U13.2, U14.1, U14.5, U14.7, U15.1, U15.2, U15.3, U15.6, U15.7, Y1.2, Y1.4

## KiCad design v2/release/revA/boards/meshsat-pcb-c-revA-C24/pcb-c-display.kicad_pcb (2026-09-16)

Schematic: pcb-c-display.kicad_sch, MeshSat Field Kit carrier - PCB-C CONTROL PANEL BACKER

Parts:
BZ1: IP67 panel-mount sounder, 5 V DC continuous, beze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; PanelSounder
C1, C2: 10u; C_0805_2012Metric; LCSC C15850
C3, C4, C14, C15, C16: 1u; C_0603_1608Metric
C5, C6: 15p NP0; C_0402_1005Metric
C7, C8, C9, C10, C11, C12, C13, C25, C29, C38: 100n; C_0603_1608Metric
C17, C18, C26, C27: 100n; C_0603_1608Metric; LCSC C14663
C19, C20, C21, C22, C23, C24: 10n; C_0603_1608Metric; LCSC C57112
C28: 4.7u; C_0805_2012Metric
C30, C31, C32, C33, C34, C35, C36, C37: 1u 25V; C_0603_1608Metric
CAM_H1, CAM_H2: M2 screw of the USB camera module (25 x 25 board,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; MountingHole_2.2mm_M2
D1: 3 mm MWARN red, sunlight viewable; LED_D3.0mm
D2: 3 mm MCAUT amber, sunlight viewable; LED_D3.0mm
D3: 3 mm TX red (RF hazard), sunlight viewable; LED_D3.0mm
D4: 3 mm SOSACT red, sunlight viewable; LED_D3.0mm
D5: 3 mm SAT green, sunlight viewable; LED_D3.0mm
D6: 3 mm MESH green, sunlight viewable; LED_D3.0mm
D7: 3 mm LTE green, sunlight viewable; LED_D3.0mm
D8: 3 mm GPS green, sunlight viewable; LED_D3.0mm
D9: 3 mm SHORE green, sunlight viewable; LED_D3.0mm
D10: 3 mm CHG white, sunlight viewable; LED_D3.0mm
D11: 3 mm MSG white, sunlight viewable; LED_D3.0mm
D12: 3 mm BAT1 amber, sunlight viewable; LED_D3.0mm
D13: 3 mm BAT2 green, sunlight viewable; LED_D3.0mm
D14: 3 mm BAT3 green, sunlight viewable; LED_D3.0mm
D15: 3 mm BAT4 green, sunlight viewable; LED_D3.0mm
D16: 3 mm BAT5 green, sunlight viewable; LED_D3.0mm
D17: BAT54 lamp-test tie; D_SOD-123; LCSC C7502705
D18: status (GPIO25); LED_0603_1608Metric
D19: SS2040FL: EPD_SW -> VGH; D_SOD-123F
D20: SS2040FL: pump clamp; D_SOD-123F
D21: SS2040FL: pump -> VGL; D_SOD-123F
FB1, FB2, FB3, FB4: ferrite 600R; L_0603_1608Metric; LCSC C1002
H1, H2, H3, H4, H5, H6, H7, H8: M3 x 6 into the face plate's self-clinching stand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; BackerScrew_M3_GND
JP1: BOOTSEL: short while powering to enter the USB bo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; SolderJumper-2_P1.3mm_Open_RoundedPad1.0x1.5mm
JP2: PANEL_ID strap (closed = variant B); SolderJumper-2_P1.3mm_Open_RoundedPad1.0x1.5mm
J_EPD: Hirose FH34SRJ-24S-0.5SH ZIF for the E2370KS0C1 f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; Hirose_FH34SRJ-24S
J_HSJ1: U-174/U headset jack 1 (Amphenol Nexus class, dra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; PanelJack_17mm
J_HSJ2: U-174/U headset jack 2 (Amphenol Nexus class, dra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; PanelJack_17mm
J_MAINSW: MAIN button lead to A22 J_MAINSW (XH2.5 at the A2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; LeadLands_1x02
J_PANEL: panel ribbon from B16 J_PANEL (IDC 2x13 SMD, unde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; IDC-Header_2x13_P2.54mm_Vertical_SMD
J_PIJ2: PI button lead: two solder lands on the underside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; LeadLands_1x02
L1: 10uH ATNR4010100MT 0.8 A (the boost inductor); L_APV_ANR4020
Q1: AO3401A P-FET high side; SOT-23; LCSC C15127
Q2, Q3, Q4: 2N7002; SOT-23; LCSC C8545
Q5: AO3401A P-FET: the e-paper's supply switch (EPD_P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; SOT-23; LCSC C15127
Q6: Si2302CDS-T1-GE3 logic-level N-FET (Vishay, SOT-2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; SOT-23; LCSC C10488
R1, R6: 1k; R_0603_1608Metric
R2, R3: 27R; R_0603_1608Metric
R4, R42: 10k; R_0603_1608Metric
R5: 1k (BOOTSEL); R_0603_1608Metric
R7, R8: 2.2k; R_0603_1608Metric
R9, R10, R11, R12, R13, R14, R15, R16: 10k; R_0603_1608Metric; LCSC C25804
R17: 2.2k; R_0603_1608Metric; LCSC C4190
R18: 47R; R_0603_1608Metric; LCSC C23182
R19, R44: 100R; R_0603_1608Metric; LCSC C22775
R20, R38, R45: 100k; R_0603_1608Metric; LCSC C25803
R21, R22, R23, R31, R36, R40: 300R; R_0603_1608Metric; LCSC C23025
R24, R25, R26, R27, R28, R29, R30, R32, R33, R34, R35: 180R; R_0603_1608Metric; LCSC C22828
R37: 1k; R_0603_1608Metric; LCSC C21190
R39, R41: 470R; R_0603_1608Metric; LCSC C23179
R43: 0.47R 1%; R_0603_1608Metric
SW_EMCON: EMCON locking toggle (closed = TX inhibit, a hard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; ToggleBody_SPDT
SW_LIGHT: LIGHTING DAY/NIGHT/BLACKOUT toggle DPDT ON-ON-ON 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; ToggleBody_DPDT
SW_MAIN: MAIN PWR 19 mm momentary, green ring (to A22 J_MA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; PanelSwitch_19mm
SW_PI: PI 16 mm recessed momentary, amber ring (PI_SHDN_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; PanelSwitch_16mm
SW_SOS: SOS locking toggle, maintained (APEM 5636ADKB-2V,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; ToggleBody_SPDT
SW_TEST: TEST/ACK 16 mm momentary, white ring; C&K ATP16-S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; PanelSwitch_16mm
SW_ZERO: ZEROIZE locking toggle, maintained (APEM 5636ADKB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; ToggleBody_SPDT
TP1: SWCLK; TestPoint_Pad_D1.5mm
TP2: SWDIO; TestPoint_Pad_D1.5mm
TP3: C_RUN; TestPoint_Pad_D1.5mm
TP4: LED_RAIL; TestPoint_Pad_D1.5mm
TP5: LED_RAIL_SW; TestPoint_Pad_D1.5mm
TP6: +5V; TestPoint_Pad_D1.5mm
TP7: +3V3; TestPoint_Pad_D1.5mm
TP8: GND; TestPoint_Pad_D1.5mm
TP9: EXP_INT; TestPoint_Pad_D1.5mm
TP10: TX_INHIBIT_n; TestPoint_Pad_D1.5mm
TP11: EMCON_HW; TestPoint_Pad_D1.5mm
TP12: ZEROIZE_HW; TestPoint_Pad_D1.5mm
TP13: SPARE1; TestPoint_Pad_D1.5mm
TP14: SPARE2; TestPoint_Pad_D1.5mm
TP15: SPARE3; TestPoint_Pad_D1.5mm
TP16: SPARE4; TestPoint_Pad_D1.5mm
TP17: SPARE5; TestPoint_Pad_D1.5mm
TP18: SPARE6; TestPoint_Pad_D1.5mm
TP19: SPARE7; TestPoint_Pad_D1.5mm
TP20: SPARE8; TestPoint_Pad_D1.5mm
TP21: SPARE9; TestPoint_Pad_D1.5mm
TP22: SPARE10; TestPoint_Pad_D1.5mm
TP23: SPARE11; TestPoint_Pad_D1.5mm
TP24: SPARE12; TestPoint_Pad_D1.5mm
TP25: EPD_BUSY; TestPoint_Pad_D1.5mm
TP26: EPD_VGH; TestPoint_Pad_D1.5mm
TP27: EPD_VGL; TestPoint_Pad_D1.5mm
TP28: HB1; TestPoint_Pad_D1.5mm
TP29: HB2; TestPoint_Pad_D1.5mm
TP30: HB3; TestPoint_Pad_D1.5mm
TP31: SLOT_EN1; TestPoint_Pad_D1.5mm
TP32: SLOT_EN2; TestPoint_Pad_D1.5mm
TP33: SLOT_EN3; TestPoint_Pad_D1.5mm
TP34: HDMI_SEL1; TestPoint_Pad_D1.5mm
TP35: HDMI_SEL2; TestPoint_Pad_D1.5mm
TP36: PI_SHDN_REQ; TestPoint_Pad_D1.5mm
TP37: PI_KILL; TestPoint_Pad_D1.5mm
TP38: SHORE_INHIBIT; TestPoint_Pad_D1.5mm
TP39: PIJ2_A; TestPoint_Pad_D1.5mm
TP40: PIJ2_B; TestPoint_Pad_D1.5mm
U1: PCA9555PW 0x22: LED sinks, light mode inputs; TSSOP-24_4.4x7.8mm_P0.65mm; LCSC C2864778
U2: PCA9555PW 0x23: LED sinks, the battery bar, lamp 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; TSSOP-24_4.4x7.8mm_P0.65mm; LCSC C2864778
U3: RP2040 panel controller (USB device on B16's slot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; QFN-56-1EP_7x7mm_P0.4mm_EP3.2x3.2mm; LCSC C2040
U4: W25Q16JVUXIQ 16 Mbit QSPI flash (USON-8: 1 CS 2 D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; Winbond_USON-8-1EP_3x2mm_P0.5mm_EP0.2x1.6mm; LCSC C2843335
U5: TLV75533PDBV 3.3 V 500 mA LDO for the controller,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; SOT-23-5
U6, U7, U8, U10, U11: USBLC6-2SC6; SOT-23-6; LCSC C7519
U9: 74LVC1G34 non-inverting buffer (2 A 4 Y): EMCON_H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; SOT-23-5
U_LIGHT: Vishay VEML7700 ambient light sensor (1 SCL 2 VDD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; Vishay_VEML7700; LCSC C504893
Y1: 12 MHz ABM8-272-T3 (3225): 1 XIN, 3 XOUT, 2 and 4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; Crystal_SMD_3225-4Pin_3.2x2.5mm; LCSC C20625731

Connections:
/+3V3: C2.1, C4.1, C7.1, C8.1, C9.1, C10.1, C11.1, C12.1, C13.1, C16.1, C17.1, C18.1, C25.1, C38.1, Q5.2 (S), R4.2, R7.2, R8.2, R9.2, R10.2, R11.2, R12.2, R13.2, R14.2, R16.2, R42.2, TP7.1, U1.2 (A1), U1.24 (VDD), U2.2 (A1), U2.21 (A0), U2.24 (VDD), U3.1 (IOVDD), U3.10 (IOVDD), U3.22 (IOVDD), U3.33 (IOVDD), U3.42 (IOVDD), U3.43 (ADC_AVDD), U3.44 (VREG_VIN), U3.48 (USB_VDD), U3.49 (IOVDD), U4.8 (+3V3), U5.5 (+3V3), U6.5 (VBUS), U7.5 (VBUS), U8.5 (VBUS), U9.5 (+3V3), U10.5 (VBUS), U11.5 (VBUS), U_LIGHT.2 (+3V3)
/+5V: BZ1.2 (-), C1.1, C3.1, J_PANEL.1, J_PANEL.2, SW_LIGHT.2, TP6.1, U5.1 (+5V), U5.3 (+5V)
/BAT1_A: D12.2 (A), R31.2
/BAT1_K: D12.1 (K), U2.7 (IO0_3)
/BAT2_A: D13.2 (A), R32.2
/BAT2_K: D13.1 (K), U2.8 (IO0_4)
/BAT3_A: D14.2 (A), R33.2
/BAT3_K: D14.1 (K), U2.9 (IO0_5)
/BAT4_A: D15.2 (A), R34.2
/BAT4_K: D15.1 (K), U2.10 (IO0_6)
/BAT5_A: D16.2 (A), R35.2
/BAT5_K: D16.1 (K), U2.11 (IO0_7)
/BOOT_J: JP1.1 (A), R5.2
/BZ_K: BZ1.1 (+), Q4.3 (D)
/CHG_A: D10.2 (A), R29.2
/CHG_K: D10.1 (K), U1.7 (IO0_3)
/C_DVDD: C14.1, C15.1, U3.23 (DVDD), U3.45 (VREG_VOUT), U3.50 (DVDD)
/C_RUN: R4.1, TP3.1, U3.26 (RUN)
/EMCON_HW: J_PANEL.8, TP11.1, U3.32 (GPIO21), U9.4 (EMCON_HW)
/EPD_BUSY: J_EPD.9 (BUSY_N), TP25.1, U3.9 (GPIO7)
/EPD_CS: J_EPD.12 (CSB), U3.7 (GPIO5)
/EPD_DC: J_EPD.11 (DC), U3.6 (GPIO4)
/EPD_GDR: J_EPD.2 (GDR), Q6.1 (G)
/EPD_PUMP: C31.2, D20.1 (K), D21.2 (A)
/EPD_PWR_n: Q5.1 (G), R42.1, U3.41 (GPIO29_A3)
/EPD_RESE: J_EPD.3 (RESE), Q6.2 (S), R43.1
/EPD_RST: J_EPD.10 (RST_N), U3.8 (GPIO6)
/EPD_SCL: J_EPD.13 (SCL), U3.4 (GPIO2)
/EPD_SDA: J_EPD.14 (SDA), U3.5 (GPIO3)
/EPD_SW: C31.1, D19.1 (K), L1.2, Q6.3 (D)
/EPD_VCC: C28.1, C29.1, J_EPD.15 (VDDIO), J_EPD.16 (VDD), L1.1, Q5.3 (D)
/EPD_VCOM: C37.1, J_EPD.24 (VCOM)
/EPD_VDDD: C34.1, J_EPD.18 (VDDD)
/EPD_VDH: C35.1, J_EPD.20 (VDH)
/EPD_VDHR: C33.1, J_EPD.5 (VDHR)
/EPD_VDL: C36.1, J_EPD.22 (VDL)
/EPD_VGH: C30.1, D19.2 (A), J_EPD.21 (VGH), TP26.1
/EPD_VGL: C32.1, D21.1 (K), J_EPD.23 (VGL), TP27.1
/EXP_INT: J_PANEL.6, TP9.1, U1.1 (~INT), U2.1 (~INT), U3.36 (GPIO24), U8.3 (I/O2), U8.4 (I/O2)
/GPS_A: D8.2 (A), R27.2
/GPS_K: D8.1 (K), U1.11 (IO0_7)
/HB1: J_PANEL.18, TP28.1, U3.13 (GPIO10)
/HB2: J_PANEL.19, TP29.1, U3.14 (GPIO11)
/HB3: J_PANEL.20, TP30.1, U3.15 (GPIO12)
/HDMI_SEL1: J_PANEL.12, TP34.1, U3.27 (GPIO16)
/HDMI_SEL2: J_PANEL.13, TP35.1, U3.28 (GPIO17)
/LED_RAIL: Q1.3 (D), R21.1, R22.1, R23.1, R24.1, R25.1, R26.1, R27.1, R28.1, R29.1, R30.1, R31.1, R32.1, R33.1, R34.1, R35.1, R36.1, R40.1, R41.1, TP4.1
/LED_RAIL_SW: Q1.2 (S), R15.1, R17.1, R39.1, SW_LIGHT.1, TP5.1
/LED_STAT: R6.1, U3.37 (GPIO25)
/LED_STAT_A: D18.2 (A), R6.2
/LIGHT_DAY_n: C22.1, R12.1, SW_LIGHT.5, U1.13 (IO1_0)
/LIGHT_NIGHT_n: C23.1, R13.1, SW_LIGHT.6, U1.14 (IO1_1)
/LTE_A: D7.2 (A), R26.2
/LTE_K: D7.1 (K), U1.10 (IO0_6)
/MAINRING_A: R39.2, SW_MAIN.3
/MAINSW_A: FB1.1, SW_MAIN.1
/MAINSW_A2: C26.1, FB1.2, J_MAINSW.1, U10.1 (I/O1), U10.6 (I/O1)
/MAINSW_B: FB2.1, SW_MAIN.2
/MAINSW_B2: C26.2, FB2.2, J_MAINSW.2, U10.3 (I/O2), U10.4 (I/O2)
/MCAUT_A: D2.2 (A), R22.2
/MCAUT_K: D2.1 (K), U1.6 (IO0_2)
/MESH_A: D6.2 (A), R25.2
/MESH_K: D6.1 (K), U1.9 (IO0_5)
/MSG_A: D11.2 (A), R30.2
/MSG_K: D11.1 (K), U2.5 (IO0_1)
/MWARN_A: D1.2 (A), R21.2
/MWARN_K: D1.1 (K), U1.5 (IO0_1)
/PANEL_ID: JP2.1 (A), R16.1, U1.15 (IO1_2)
/PANEL_PWM: R19.1, U3.11 (GPIO8)
/PIJ2_A: FB3.1, SW_PI.1, TP39.1
/PIJ2_A2: C27.1, FB3.2, J_PIJ2.1, U11.1 (I/O1), U11.6 (I/O1)
/PIJ2_B: FB4.1, SW_PI.2, TP40.1
/PIJ2_B2: C27.2, FB4.2, J_PIJ2.2, U11.3 (I/O2), U11.4 (I/O2)
/PIRING_A: R40.2, SW_PI.3
/PIRING_K: SW_PI.4, U2.6 (IO0_2)
/PI_KILL: J_PANEL.25, TP37.1, U3.30 (GPIO19)
/PI_SHDN_REQ: J_PANEL.24, TP36.1, U3.29 (GPIO18)
/PWM1: R44.1, U3.12 (GPIO9)
/Q1_G: Q1.1 (G), R17.2, R18.1
/Q2_D: Q2.3 (D), R18.2
/Q2_G: Q2.1 (G), R19.2, R20.1
/Q3_G: Q3.1 (G), R37.2, R38.1
/Q4_G: Q4.1 (G), R44.2, R45.1
/QSPI_D0: U3.53 (QSPI_SD0), U4.5 (QSPI_D0)
/QSPI_D1: U3.55 (QSPI_SD1), U4.2 (QSPI_D1)
/QSPI_D2: U3.54 (QSPI_SD2), U4.3 (QSPI_D2)
/QSPI_D3: U3.51 (QSPI_SD3), U4.7 (QSPI_D3)
/QSPI_SCLK: U3.52 (QSPI_SCLK), U4.6 (QSPI_SCLK)
/QSPI_SS: R5.1, U3.56 (QSPI_SS_N), U4.1 (QSPI_SS)
/RAIL_SENSE: R15.2, U3.38 (GPIO26_A0)
/SAT_A: D5.2 (A), R24.2
/SAT_K: D5.1 (K), U1.8 (IO0_4)
/SCL: J_PANEL.5, R8.1, U1.22 (SCL), U2.22 (SCL), U3.3 (GPIO1), U7.3 (I/O2), U7.4 (I/O2), U_LIGHT.1 (SCL)
/SDA: J_PANEL.4, R7.1, U1.23 (SDA), U2.23 (SDA), U3.2 (GPIO0), U7.1 (I/O1), U7.6 (I/O1), U_LIGHT.4 (SDA)
/SHORE_A: D9.2 (A), R28.2
/SHORE_INHIBIT: J_PANEL.26, TP38.1, U3.31 (GPIO20)
/SHORE_K: D9.1 (K), U2.4 (IO0_0)
/SLOT_EN1: J_PANEL.21, TP31.1, U3.16 (GPIO13)
/SLOT_EN2: J_PANEL.22, TP32.1, U3.17 (GPIO14)
/SLOT_EN3: J_PANEL.23, TP33.1, U3.18 (GPIO15)
/SOSACT_A: D4.2 (A), R23.2
/SOSACT_K: D4.1 (K), U1.4 (IO0_0)
/SOS_SW: C19.1, R9.1, SW_SOS.1, U3.40 (GPIO28_A2)
/SPARE1: TP13.1, U1.16 (IO1_3)
/SPARE2: TP14.1, U1.17 (IO1_4)
/SPARE3: TP15.1, U1.18 (IO1_5)
/SPARE4: TP16.1, U1.19 (IO1_6)
/SPARE5: TP17.1, U1.20 (IO1_7)
/SPARE6: TP18.1, U2.14 (IO1_1)
/SPARE7: TP19.1, U2.15 (IO1_2)
/SPARE8: TP20.1, U2.16 (IO1_3)
/SPARE9: TP21.1, U2.17 (IO1_4)
/SPARE10: TP22.1, U2.18 (IO1_5)
/SPARE11: TP23.1, U2.19 (IO1_6)
/SPARE12: TP24.1, U2.20 (IO1_7)
/SWCLK: TP1.1, U3.24 (SWCLK)
/SWDIO: TP2.1, U3.25 (SWD)
/TESTRING_A: R41.2, SW_TEST.3
/TEST_SW: C21.1, R11.1, SW_TEST.1, U3.39 (GPIO27_A1)
/TR_APRS: J_PANEL.7, R37.1, U3.35 (GPIO23), U8.1 (I/O1), U8.6 (I/O1)
/TX_A: D3.2 (A), R36.2
/TX_INHIBIT_n: C24.1, J_PANEL.11, R14.1, SW_EMCON.1, TP10.1, U9.2 (TX_INHIBIT_n)
/TX_K: D3.1 (K), D17.2 (A), Q3.3 (D)
/TX_LAMPTEST: D17.1 (K), U2.13 (IO1_0)
/USB_DM_R: R3.1, U3.46 (USB_DM)
/USB_DP_R: R2.1, U3.47 (USB_DP)
/USB_PNL_N: J_PANEL.16, R3.2, U6.3 (I/O2), U6.4 (I/O2)
/USB_PNL_P: J_PANEL.15, R2.2, U6.1 (I/O1), U6.6 (I/O1)
/XIN: C5.1, U3.20 (XIN), Y1.1
/XOUT: C6.1, R1.2, Y1.3
/XOUT_R: R1.1, U3.21 (XOUT)
/ZEROIZE_HW: C20.1, J_PANEL.10, R10.1, SW_ZERO.1, TP12.1, U3.34 (GPIO22)
GND: C1.2, C2.2, C3.2, C4.2, C5.2, C6.2, C7.2, C8.2, C9.2, C10.2, C11.2, C12.2, C13.2, C14.2, C15.2, C16.2, C17.2, C18.2, C19.2, C20.2, C21.2, C22.2, C23.2, C24.2, C25.2, C28.2, C29.2, C30.2, C32.2, C33.2, C34.2, C35.2, C36.2, C37.2, C38.2, D18.1 (K), D20.2 (A), H1.1, H2.1, H3.1, H4.1, H5.1, H6.1, H7.1, H8.1, JP1.2 (B), JP2.2 (B), J_EPD.8 (BS), J_EPD.17 (VSS), J_EPD.25 (SHIELD), J_EPD.26 (SHIELD), J_PANEL.3, J_PANEL.9, J_PANEL.14, J_PANEL.17, Q2.2 (S), Q3.2 (S), Q4.2 (S), R20.2, R38.2, R43.2, R45.2, SW_EMCON.2, SW_LIGHT.4, SW_MAIN.4, SW_SOS.2, SW_TEST.2, SW_TEST.4, SW_ZERO.2, TP8.1, U1.3 (A2), U1.12 (VSS), U1.21 (A0), U2.3 (A2), U2.12 (VSS), U3.19 (TESTEN), U3.57 (GND), U4.4 (GND), U4.9 (GND), U5.2 (GND), U6.2 (GND), U7.2 (GND), U8.2 (GND), U9.3 (GND), U10.2 (GND), U11.2 (GND), U_LIGHT.3 (GND), Y1.2 (G), Y1.4 (G)

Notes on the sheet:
PCB-C CONTROL PANEL BACKER C24
RIBBON FROM B16, 5 V, 3.3 V LDO, USB AND BUS ESD, FLAGS | RP2040 PANEL CONTROLLER, FLASH, CRYSTAL, BOOTSEL, BUS PULL-UPS
RIBBON FROM B16, 5 V, 3.3 V LDO, USB AND BUS ESD, FLAGS
RP2040 PANEL CONTROLLER, FLASH, CRYSTAL, BOOTSEL, BUS PULL-UPS
page 1 of 5 MeshSat field kit V2, CERN-OHL-S-2.0 PROTOTYPE, nothing built 2026-09-16
panel ribbon from B16 J_PANEL
TLV75533PDBV 3.3 V 500 mA LDO for..
RP2040 panel controller
status
BOOTSEL
p2,5
p2,4,5
p2,3,4
p3,4
p4,5
p2,4
RP2040 PANEL CONTROLLER, FLASH, CRYSTAL, BOOTSEL, BUS PULL-UPS | EXPANDERS 0x22 / 0x23, MODE INPUTS, EMCON INVERTER, STRAPS | LED RAIL, INDICATORS, TX LAMP, SWITCHES
RP2040 PANEL CONTROLLER, FLASH, CRYSTAL, BOOTSEL, BUS PULL-UPS (continued)
EXPANDERS 0x22 / 0x23, MODE INPUTS, EMCON INVERTER, STRAPS
LED RAIL, INDICATORS, TX LAMP, SWITCHES AND LEADS
page 2 of 5 MeshSat field kit V2, CERN-OHL-S-2.0 PROTOTYPE, nothing built 2026-09-16
W25Q16JVUXIQ 16 Mbit QSPI flash
12 MHz ABM8-272-T3
PCA9555PW 0x22
PANEL_ID strap
PCA9555PW 0x23
74LVC1G34 non-inverting buffer
LIGHTING DAY/NIGHT/BLACKOUT toggle..
p1,5
p1,4,5
p1,4
p1,3,4
LED RAIL, INDICATORS, TX LAMP, SWITCHES AND LEADS (continued)
page 3 of 5 MeshSat field kit V2, CERN-OHL-S-2.0 PROTOTYPE, nothing built 2026-09-16
3 mm MWARN red
3 mm MCAUT amber
3 mm SOSACT red
3 mm SAT green
3 mm MESH green
3 mm LTE green

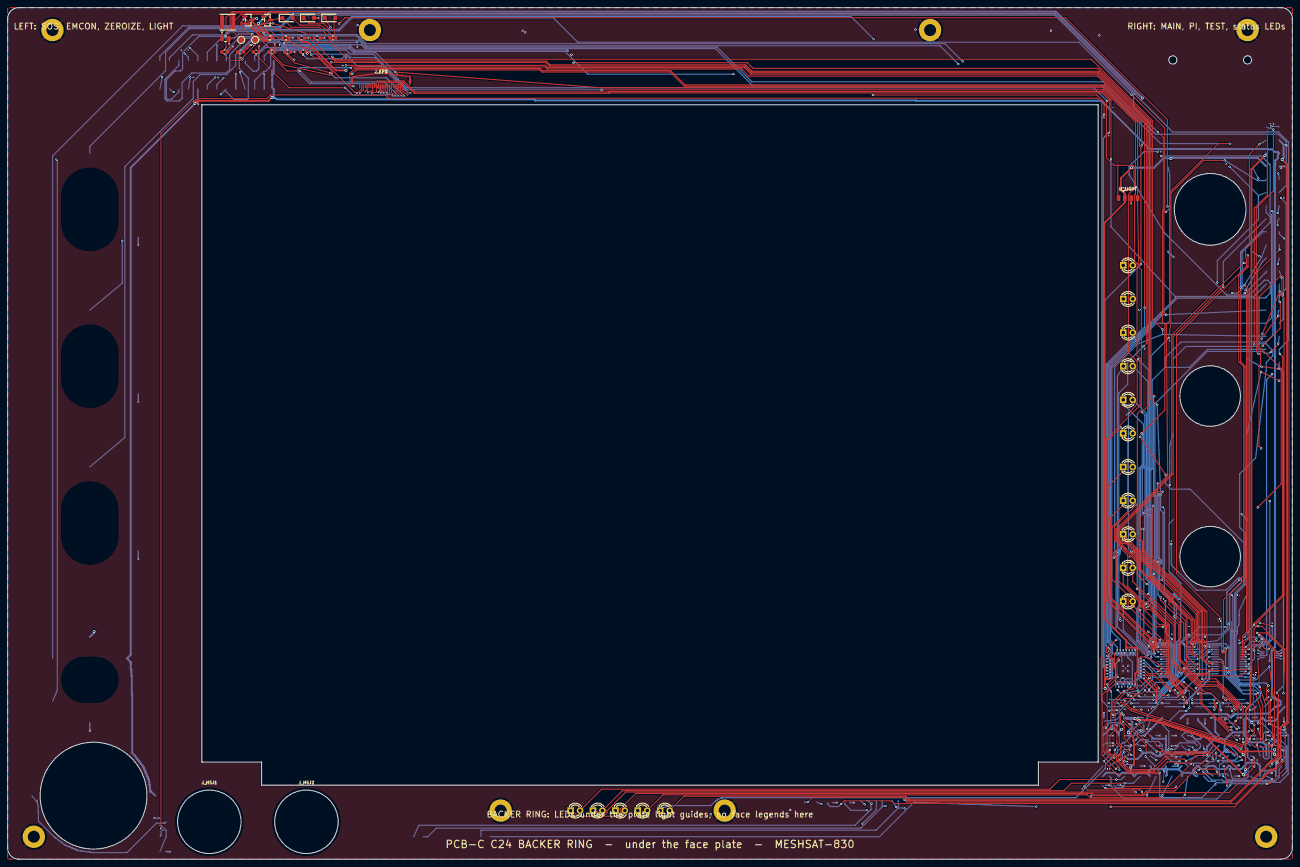
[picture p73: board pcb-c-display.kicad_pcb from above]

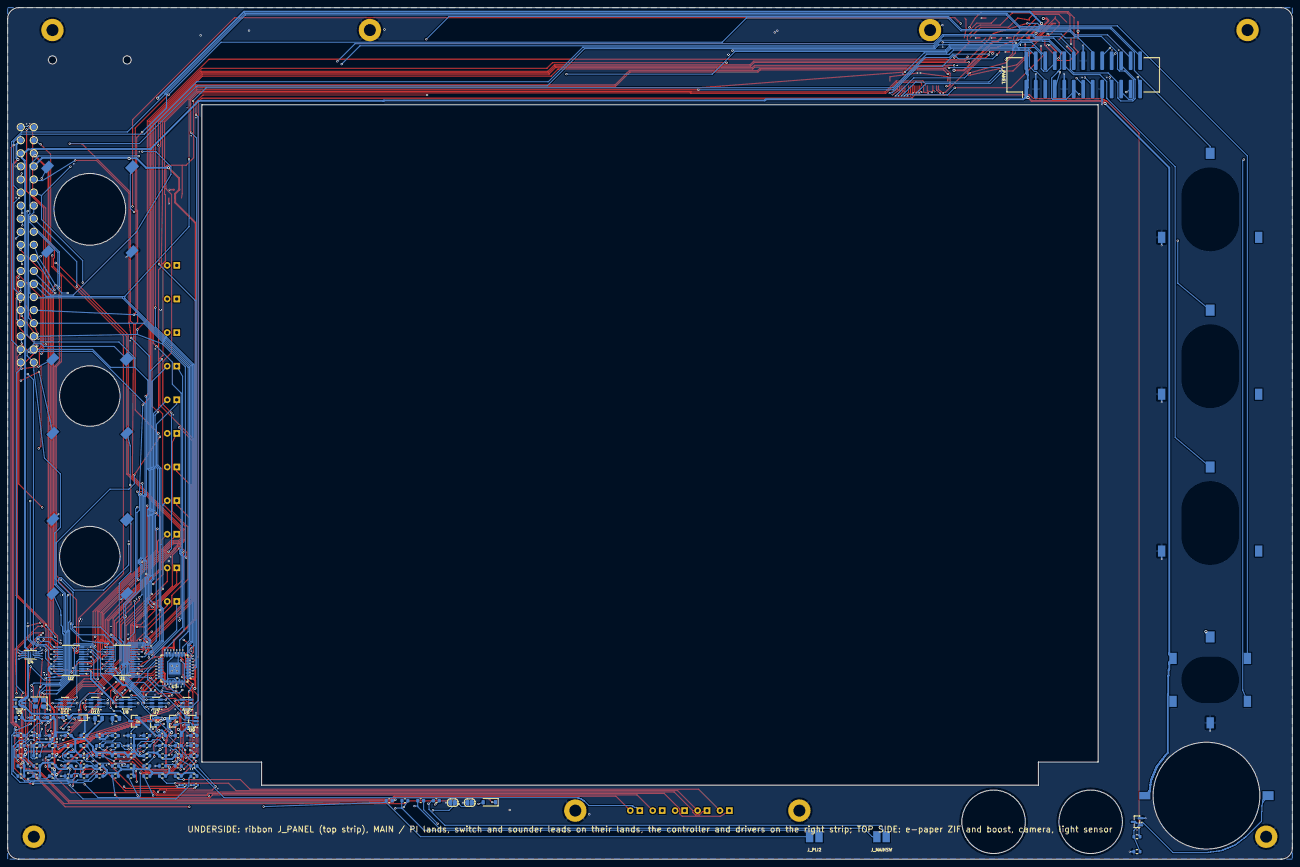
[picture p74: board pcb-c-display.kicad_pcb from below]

Board: 4 copper layers, 344.0 x 228.0 mm, 194 parts (135 on the bottom side), 133 nets.

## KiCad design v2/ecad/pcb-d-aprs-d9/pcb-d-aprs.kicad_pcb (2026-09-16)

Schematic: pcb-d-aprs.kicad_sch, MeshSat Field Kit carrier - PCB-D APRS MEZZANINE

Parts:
C1, C2, C5: 47u 6.3V X5R 1210; C_1210_3225Metric
C3, C9, C17, C24, C25, C33, C40: 10u; C_0805_2012Metric
C4, C6, C11, C15, C16, C39, C49, C50, C51, C52, C53, C54, C55, C56, C57, C62, C63: 100n; C_0603_1608Metric
C7, C8, C12, C18, C19, C20, C21, C22, C23, C28, C29, C30, C31, C32, C34, C35, C36, C37, C38, C41, C42, C46, C47, C48: 1u; C_0603_1608Metric
C10: 4.7u; C_0805_2012Metric
C13, C14: 27p NP0; C_0402_1005Metric
C26, C27: 18p NP0; C_0402_1005Metric
C43: 100p NP0; C_0402_1005Metric
C44, C45: 1n NP0; C_0402_1005Metric
C58, C60: 22p 500V NP0 1206; C_1206_3216Metric
C59: 39p 500V NP0 1206; C_1206_3216Metric
C61: 4.7n; C_0402_1005Metric
D1: SMBJ5.0A; D_SMB
D2: 1N4148W coil flyback; D_SOD-123
FB1: 600R 2A ferrite (the exciter's 1 A transmit pulse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; L_0805_2012Metric
JP1: electret bias headset 1 (close for an electret mi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; SolderJumper-2_P1.3mm_Open_RoundedPad1.0x1.5mm
JP2: electret bias headset 2; SolderJumper-2_P1.3mm_Open_RoundedPad1.0x1.5mm
J_ANT: SMA jack: antenna pigtail to A22's VHF jack J_RF1; SMA_Amphenol_132134_Vertical; LCSC C3174425
J_HARN1: A22 mezzanine harness J_MEZZ1 (IDC 2x8): USB pair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; IDC-Header_2x08_P2.54mm_Vertical_NarrowPad
J_HS1: JST-PH 1x5 socket: headset 1, SPK GND MIC GND PTT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; JST_PH_B5B-PH-K_1x05_P2.00mm_Vertical; LCSC C157993
J_HS2: JST-PH 1x5 socket: headset 2, SPK GND MIC GND PTT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; JST_PH_B5B-PH-K_1x05_P2.00mm_Vertical; LCSC C157993
J_PAIN: U.FL socket: PA drive (coax to the RA30H1317M1 in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; U.FL_Hirose_U.FL-R-SMT-1_Vertical; LCSC C88373
J_PAOUT: SMA jack: PA output (coax from the RA30H1317M1 ou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; SMA_Amphenol_132134_Vertical; LCSC C3174425
J_PWR1: JST-VH socket, 10 A: 5 V from A22 J_MEZZ_PWR1 (be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; JST_VH_B2P-VH_1x02_P3.96mm_Vertical; LCSC C274411
J_USB3: JST-PH 1x4 socket: spare hub port 3, 5V D- D+ GND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; JST_PH_B4B-PH-K_1x04_P2.00mm_Vertical; LCSC C131334
J_VGG: JST-PH 1x2 socket: PA gate bias, VGG GND (the lea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; JST_PH_B2B-PH-K_1x02_P2.00mm_Vertical; LCSC C5251182
K1: Omron G6K-2F-Y 5 VDC DPDT signal relay, T/R; Relay_DPDT_Omron_G6K-2F-Y
L1: 68nH 0805 (LPF, 145 MHz 5th order; values to be v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; L_0805_2012Metric
L2: 68nH 0805 (LPF); L_0805_2012Metric
LED1: green power; LED_0603_1608Metric; LCSC C12624
LED2: amber record; LED_0603_1608Metric; LCSC C2287
LED3: green playback; LED_0603_1608Metric; LCSC C12624
LED4: red transmit; LED_0603_1608Metric; LCSC C2286
LED5: amber PA keyed; LED_0603_1608Metric; LCSC C2287
LED6: green receive (AUDIO_ON low); LED_0603_1608Metric; LCSC C12624
Q1: 2N7002 PA_EN -> H/L low (never tie H/L high); SOT-23; LCSC C8545
Q2: 2N7002 relay coil; SOT-23; LCSC C8545
Q3, Q4, Q5, Q6, Q7, Q8, Q9: 2N7002; SOT-23; LCSC C8545
R1, R43, R44, R51: 2.2k; R_0603_1608Metric
R2, R3, R34, R53: 100k; R_0603_1608Metric
R4, R29, R30, R49, R50, R52: 1k; R_0603_1608Metric
R5, R9, R10, R31, R32, R35, R36, R37, R38, R39, R45, R46, R47, R66, R67, R68, R69, R70, R71, R72, R73, R74, R75, R76, R77, R78, R79: 10k; R_0603_1608Metric
R6, R7, R12, R13, R16, R17, R20, R21: 22; R_0603_1608Metric
R8, R11, R28: 1.5k; R_0603_1608Metric
R14, R15, R18, R19, R22, R23, R24, R25: 15k; R_0603_1608Metric
R26, R27: 33; R_0603_1608Metric
R33, R40, R41: 4.7k; R_0603_1608Metric
R42: 220k; R_0603_1608Metric
R48: 100; R_0603_1608Metric
R54, R56: 27 1% 2010; R_2010_5025Metric
R55: 36 1% 2010; R_2010_5025Metric
TP1: AF_OUT; TestPoint_Pad_D1.5mm
TP2: MIC_SUM; TestPoint_Pad_D1.5mm
TP3: KEY; TestPoint_Pad_D1.5mm
TP4: PA_KEY; TestPoint_Pad_D1.5mm
TP5: +3V3_D8; TestPoint_Pad_D1.5mm
TP6: +5V_D8; TestPoint_Pad_D1.5mm
TP7: VGG_SW; TestPoint_Pad_D1.5mm
TP8: RX_MIX; TestPoint_Pad_D1.5mm
TP9: ZEROIZE_HW; TestPoint_Pad_D1.5mm
TP10: AB_SPARE; TestPoint_Pad_D1.5mm
TP11: SA_TXD; TestPoint_Pad_D1.5mm
TP12: SA_RXD; TestPoint_Pad_D1.5mm
TP13: PTT_SW_n; TestPoint_Pad_D1.5mm
TP14: SA_PD; TestPoint_Pad_D1.5mm
TP15: TX_INHIBIT_n; TestPoint_Pad_D1.5mm
TP16: PA_EN; TestPoint_Pad_D1.5mm
TP17: EXP_SPARE1; TestPoint_Pad_D1.5mm
TP18: EXP_SPARE2; TestPoint_Pad_D1.5mm
TP19: EXP_SPARE3; TestPoint_Pad_D1.5mm
TP20: EXP_SPARE4; TestPoint_Pad_D1.5mm
TP21: EXP_SPARE5; TestPoint_Pad_D1.5mm
TP22: EXP_SPARE6; TestPoint_Pad_D1.5mm
TP23: EXP_SPARE7; TestPoint_Pad_D1.5mm
TP24: EXP_SPARE8; TestPoint_Pad_D1.5mm
U1: TLV75533PDBV 3.3 V 500 mA LDO (1 IN 2 GND 3 EN 4 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; SOT-23-5
U2: NiceRF SA868 VHF 2 W exciter, bench-fitted (caste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; NiceRF_SA868
U3: CP2102N-A02-GQFN28 USB-UART bridge (SAU); QFN-28-1EP_5x5mm_P0.5mm_EP3.35x3.35mm; LCSC C964632
U4: TUSB2046BI four-port USB 2.0 full-speed hub (LQFP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; LQFP-32_7x7mm_P0.8mm
U5: USBLC6-2SC6; SOT-23-6; LCSC C7519
U6: TI PCM2912A USB audio codec (TQFP-32): mono input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; TQFP-32_7x7mm_P0.8mm
U7: TI TPA6132A2 headphone amplifier (QFN-16), receiv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; QFN-16-1EP_3x3mm_P0.5mm_EP1.75x1.75mm
U8: TLV9062IDGK dual op amp (1 OUT1 2 IN1- 3 IN1+ 4 V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; VSSOP-8_3x3mm_P0.65mm
U9: 74LVC1G08 AND (1 A 2 B 3 GND 4 Y 5 VCC): both hea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; SOT-23-5
U10: 74LVC1G08 AND: headsets AND software PTT (RTS); SOT-23-5
U11: 74LVC1G04 inverter (2 A 4 Y): PTT_ANY; SOT-23-5
U12: 74LVC1G08 AND: KEY = PTT_ANY AND TX_INHIBIT_n (th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; SOT-23-5
U13: 74LVC1G04 inverter: KEY -> SA868 PTT (low = trans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; SOT-23-5
U14: 74LVC1G08 AND: PA_KEY = KEY AND PA_EN (A22's PA r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; SOT-23-5
U15: TPS22810DRV; WSON-6-1EP_2x2mm_P0.65mm_EP1x1.6mm
U16: PCA9555PW 0x26: COS, PTT states, KEY, PA_KEY in; 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; TSSOP-24_4.4x7.8mm_P0.65mm
Y1: 6 MHz 3225 (CL 20 pF; C1 = C2 = 27 pF and Rd 1.5k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; Crystal_SMD_3225-4Pin_3.2x2.5mm
Y2: 6 MHz 3225 (codec clock; 18 pF loads, to confirm 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; Crystal_SMD_3225-4Pin_3.2x2.5mm

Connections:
/+3V3: C63.1, J_HARN1.13, R67.2, R69.2, R71.2, R73.2, R75.2, R77.2, R79.2, U16.2 (A1), U16.3 (A2), U16.24 (VDD)
/+3V3_D8: C8.1, C9.1, C15.1, C16.1, C17.1, C51.1, C52.1, C53.1, C54.1, C55.1, C56.1, Q3.1 (G), Q4.1 (G), Q5.1 (G), Q6.1 (G), Q7.1 (G), Q8.1 (G), Q9.1 (G), R1.1, R5.2, R8.2, R9.2, R10.2, R29.1, R30.1, R51.1, R66.2, R68.2, R70.2, R72.2, R74.2, R76.2, R78.2, TP5.1, U1.5 (+3V3_D8), U4.3 (VCC), U4.6 (EEDATA/GANGED), U4.25 (VCC), U4.26 (EXTMEM), U7.6 (G0), U9.5 (+3V3_D8), U10.5 (+3V3_D8), U11.5 (+3V3_D8), U12.5 (+3V3_D8), U13.5 (+3V3_D8), U14.5 (+3V3_D8)
/+5V_D8: C1.1, C2.1, C3.1, C4.1, C7.1, C18.1, C32.1, C33.1, C39.1, C57.1, D1.2 (A2), D2.1 (K), FB1.1, J_PWR1.1, J_USB3.1, K1.1, R38.1, R43.2, R44.2, TP6.1, U1.1 (+5V_D8), U1.3 (+5V_D8), U3.7 (VREGIN), U3.8 (VBUS), U5.5 (VBUS), U6.2 (VBUS), U7.14 (VDD), U8.8 (+5V_D8), U15.6 (VIN)
/+5V_SA: C5.1, C6.1, FB1.2, U2.8 (VBAT)
/AB_SPARE: J_HARN1.16, TP10.1
/AF_DIV: C28.1, R31.2, R32.1
/AF_OUT: R31.1, R35.1, TP1.1, U2.3 (AF_OUT)
/AMP_CPN: C30.2, U7.9 (CPN)
/AMP_CPP: C30.1, U7.11 (CPP)
/AMP_EN: Q9.2 (S), R78.1, U7.13 (EN)
/AMP_HPVDD: C31.1, U7.12 (HPVDD)
/AMP_HPVSS: C29.1, U7.8 (HPVSS)
/AMP_INL_N: C37.1, U7.1 (INL-)
/AMP_INL_P: C35.2, U7.2 (INL+)
/AMP_INR_N: C38.1, U7.4 (INR-)
/AMP_INR_P: C36.2, U7.3 (INR+)
/EXP_INT: J_HARN1.12, U16.1 (~INT)
/EXP_SPARE1: TP17.1, U16.13 (IO1_0)
/EXP_SPARE2: TP18.1, U16.14 (IO1_1)
/EXP_SPARE3: TP19.1, U16.15 (IO1_2)
/EXP_SPARE4: TP20.1, U16.16 (IO1_3)
/EXP_SPARE5: TP21.1, U16.17 (IO1_4)
/EXP_SPARE6: TP22.1, U16.18 (IO1_5)
/EXP_SPARE7: TP23.1, U16.19 (IO1_6)
/EXP_SPARE8: TP24.1, U16.20 (IO1_7)
/HS1_BIAS_R: JP1.2 (B), R43.1
/HS1_MIC: C41.1, C44.1, JP1.1 (A), J_HS1.3
/HS1_MIC_AC: C41.2, R40.1
/HS1_SPK: J_HS1.1, U7.16 (OUTL)
/HS2_BIAS_R: JP2.2 (B), R44.1
/HS2_MIC: C42.1, C45.1, JP2.1 (A), J_HS2.3
/HS2_MIC_AC: C42.2, R41.1
/HS2_SPK: J_HS2.1, U7.5 (OUTR)
/HUB_DM0: R7.2, U4.2 (DM0)
/HUB_DM1: R13.1, U4.11 (DM1)
/HUB_DM2: R17.1, U4.15 (DM2)
/HUB_DM3: R21.1, U4.19 (DM3)
/HUB_DM4: R25.1, U4.23 (DM4)
/HUB_DP0: R6.2, R8.1, U4.1 (DP0)
/HUB_DP1: R12.1, U4.12 (DP1)
/HUB_DP2: R16.1, U4.16 (DP2)
/HUB_DP3: R20.1, U4.20 (DP3)
/HUB_DP4: R24.1, U4.24 (DP4)
/HUB_OVRCUR_n: R9.1, U4.10 (OVRCUR1_n), U4.14 (OVRCUR2_n), U4.18 (OVRCUR3_n), U4.22 (OVRCUR4_n)
/HUB_RST_n: C12.1, R10.1, U4.4 (RESET_n)
/HUB_XTAL1: C13.1, U4.30 (XTAL1), Y1.1
/HUB_XTAL2: R11.2, U4.29 (XTAL2)
/HUB_XTAL2R: C14.1, R11.1, Y1.3
/KEY: Q6.2 (S), R48.1, R49.1, R72.1, TP3.1, U12.4 (KEY), U13.2 (KEY), U14.1 (KEY)
/LED_PA_A: LED5.2 (A), R50.2
/LED_PLAY_A: LED3.2 (A), R30.2
/LED_PLAY_K: LED3.1 (K), U6.32 (PLAY)
/LED_PWR_A: LED1.2 (A), R1.2
/LED_REC_A: LED2.2 (A), R29.2
/LED_REC_K: LED2.1 (K), U6.31 (REC)
/LED_RX_A: LED6.2 (A), R51.2
/LED_TX_A: LED4.2 (A), R49.2
/MICAMP_AC: C46.2, R45.1
/MICAMP_IN_N: C43.2, R40.2, R41.2, R42.2, U8.2 (MICAMP_IN_N)
/MICAMP_OUT: C43.1, C46.1, R42.1, U8.1 (MICAMP_OUT)
/MIC_IN: C48.2, U2.18 (MIC_IN)
/MIC_SUM: C48.1, R45.2, R46.2, R47.1, TP2.1
/MMUTE: R33.2, R34.1, U6.30 (MMUTE)
/OPB_OUT: U8.6 (OPB_OUT), U8.7 (OPB_OUT)
/PA_EN: J_HARN1.9, Q1.1 (G), R3.1, TP16.1, U14.2 (PA_EN)
/PA_KEY: Q7.2 (S), R50.1, R52.1, R74.1, TP4.1, U14.4 (PA_KEY), U15.5 (EN/UVLO)
/PCM_L_AC: C34.2, R36.1
/PCM_R_AC: C47.2, R46.1
/PCM_VCCA: C20.1, U6.15 (VCCA)
/PCM_VCCL: C21.1, U6.19 (VCCL)
/PCM_VCCP: C23.1, U6.26 (VCCP)
/PCM_VCCR: C22.1, U6.21 (VCCR)
/PCM_VCOM1: C24.1, U6.11 (VCOM1)
/PCM_VCOM2: C25.1, U6.12 (VCOM2)
/PCM_VDD: C19.1, R28.2, U6.5 (VDD), U6.27 (TEST1)
/PCM_VIN: C28.2, U6.16 (VIN)
/PCM_VOUTL: C34.1, U6.18 (VOUTL)
/PCM_VOUTR: C47.1, U6.22 (VOUTR)
/PCM_XTI: C26.1, U6.8 (XTI), Y2.1
/PCM_XTO: C27.1, U6.7 (XTO), Y2.3
/PTT_ANY: U11.4 (PTT_ANY), U12.1 (PTT_ANY)
/PTT_ANY_n: U10.4 (PTT_ANY_n), U11.2 (PTT_ANY_n)
/PTT_HS1_n: C49.1, J_HS1.5, Q4.2 (S), R68.1, U9.1 (PTT_HS1_n)
/PTT_HS2_n: C50.1, J_HS2.5, Q5.2 (S), R70.1, U9.2 (PTT_HS2_n)
/PTT_HS_n: U9.4 (PTT_HS_n), U10.1 (PTT_HS_n)
/PTT_SW_n: R5.1, TP13.1, U3.24 (RTS), U10.2 (PTT_SW_n)
/RF_ANT: J_ANT.1 (In), K1.6
/RF_DRV: J_PAIN.1 (In), R56.2
/RF_LPF_M: C59.1, L1.2, L2.1
/RF_LPF_OUT: C60.1, K1.5, L2.2
/RF_PAD_IN: K1.4, R54.1
/RF_PAD_M: R54.2, R55.1, R56.1
/RF_PAOUT: C58.1, J_PAOUT.1 (In), L1.1
/RF_RX: K1.2, K1.7
/RF_SA: K1.3, U2.12 (ANT)
/RLY_DRV: Q2.1 (G), R52.2, R53.1
/RLY_K: D2.2 (A), K1.8, Q2.3 (D)
/RX_MIX: C35.1, C36.1, R35.2, R36.2, R37.1, TP8.1
/SAU_3V3: C10.1, C11.1, R4.2, U3.6 (VDD)
/SAU_RST: R4.1, U3.9 (RSTb)
/SA_AUDIO_ON_n: LED6.1 (K), Q3.2 (S), R66.1, U2.1 (AUDIO_ON_n)
/SA_HL: Q1.3 (D), U2.7 (H/L)
/SA_PD: Q8.2 (S), R76.1, TP14.1, U2.6 (PD)
/SA_PTT_n: U2.5 (PTT_n), U13.4 (SA_PTT_n)
/SA_RXD: TP12.1, U2.16 (RXD), U3.26 (TXD)
/SA_TXD: TP11.1, U2.17 (TXD), U3.25 (RXD)
/SCL: J_HARN1.11, U16.22 (SCL)
/SDA: J_HARN1.10, U16.23 (SDA)
/TR_APRS: J_HARN1.7, R48.2
/TX_INHIBIT_n: J_HARN1.8, R2.1, TP15.1, U12.2 (TX_INHIBIT_n)
/USB1_N: R13.2, R15.1, R27.1
/USB1_NR: R27.2, U6.3 (D-)
/USB1_P: R12.2, R14.1, R26.1
/USB1_PR: R26.2, R28.1, U6.4 (D+)
/USB2_N: R17.2, R19.1, U3.5 (D-)
/USB2_P: R16.2, R18.1, U3.4 (D+)
/USB3_N: J_USB3.2, R21.2, R23.1
/USB3_P: J_USB3.3, R20.2, R22.1
/USB_D8_N: J_HARN1.2, R7.1, U5.3 (I/O2), U5.4 (I/O2)
/USB_D8_P: J_HARN1.1, R6.1, U5.1 (I/O1), U5.6 (I/O1)
/VGG_CT: C61.1, U15.3 (CT)
/VGG_SW: C62.1, J_VGG.1, TP7.1, U15.1 (VOUT)
/VREF: C40.1, R38.2, R39.1, U8.3 (VREF), U8.5 (VREF)
/X_AMP_EN: Q9.3 (D), R79.1, U16.10 (IO0_6)
/X_COS_n: Q3.3 (D), R67.1, U16.4 (IO0_0)
/X_KEY: Q6.3 (D), R73.1, U16.7 (IO0_3)
/X_MMUTE: R33.1, U16.11 (IO0_7)
/X_PA_KEY: Q7.3 (D), R75.1, U16.8 (IO0_4)
/X_PTT_HS1_n: Q4.3 (D), R69.1, U16.5 (IO0_1)
/X_PTT_HS2_n: Q5.3 (D), R71.1, U16.6 (IO0_2)
/X_SA_PD: Q8.3 (D), R77.1, U16.9 (IO0_5)
/ZEROIZE_HW: J_HARN1.15, TP9.1
GND: C1.2, C2.2, C3.2, C4.2, C5.2, C6.2, C7.2, C8.2, C9.2, C10.2, C11.2, C12.2, C13.2, C14.2, C15.2, C16.2, C17.2, C18.2, C19.2, C20.2, C21.2, C22.2, C23.2, C24.2, C25.2, C26.2, C27.2, C29.2, C31.2, C32.2, C33.2, C37.2, C38.2, C39.2, C40.2, C44.2, C45.2, C49.2, C50.2, C51.2, C52.2, C53.2, C54.2, C55.2, C56.2, C57.2, C58.2, C59.2, C60.2, C61.2, C62.2, C63.2, D1.1 (A1), J_ANT.2 (Ext), J_HARN1.3, J_HARN1.4, J_HARN1.5, J_HARN1.6, J_HARN1.14, J_HS1.2, J_HS1.4, J_HS2.2, J_HS2.4, J_PAIN.2 (Ext), J_PAOUT.2 (Ext), J_PWR1.2, J_USB3.4, J_VGG.2, LED1.1 (K), LED4.1 (K), LED5.1 (K), Q1.2 (S), Q2.2 (S), R2.2, R3.2, R14.2, R15.2, R18.2, R19.2, R22.2, R23.2, R24.2, R25.2, R32.2, R34.2, R37.2, R39.2, R47.2, R53.2, R55.2, U1.2 (GND), U2.9 (GND), U2.10 (GND), U3.3 (GND), U3.29 (GND), U4.7 (GND), U4.8 (BUSPWR), U4.27 (TSTPLL/48MCLK), U4.28 (GND), U4.31 (TSTMODE), U5.2 (GND), U6.1 (BGND), U6.6 (DGND), U6.13 (AGND), U6.20 (HGND), U6.23 (MAMP), U6.24 (POWER), U6.25 (PGND), U6.28 (TEST0), U7.7 (G1), U7.10 (PGND), U7.15 (SGND), U7.17 (PAD), U8.4 (GND), U9.3 (GND), U10.3 (GND), U11.3 (GND), U12.3 (GND), U13.3 (GND), U14.3 (GND), U15.4 (GND), U15.7 (GND), U16.12 (VSS), U16.21 (A0), Y1.2 (G), Y1.4 (G), Y2.2 (G), Y2.4 (G)

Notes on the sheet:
PCB-D APRS MEZZANINE D12
HARNESS, 5 V ENTRY, 3.3 V LDO, EXCITER SUPPLY | SA868 EXCITER, UART BRIDGE, T/R RELAY, 10 dB PAD, LPF, PA LEADS, GATE BIAS SWITCH
HARNESS, 5 V ENTRY, 3.3 V LDO, EXCITER SUPPLY
SA868 EXCITER, UART BRIDGE, T/R RELAY, 10 dB PAD, LPF, PA LEADS, GATE BIAS SWITCH
page 1 of 5 MeshSat field kit V2, CERN-OHL-S-2.0 PROTOTYPE, nothing built 2026-09-16
A22 mezzanine harness J_MEZZ1
JST-VH socket
47u 6.3V
600R 2A
TLV75533PDBV 3.3 V 500 mA LDO
NiceRF SA868 VHF 2 W exciter
2N7002 PA_EN -> H/L low
CP2102N-A02-GQFN28 USB-UART bridge
Omron G6K-2F-Y 5 VDC DPDT signal r..
27 1%
68nH 0805
U.FL socket
SMA jack
22p 500V
39p 500V
p4,5
p3,5
SA868 EXCITER, UART BRIDGE, T/R RELAY, 10 dB PAD, LPF, PA LEADS, GATE BIAS SWITCH | USB HUB TUSB2046B, PORT TERMINATIONS, SPARE PORT
SA868 EXCITER, UART BRIDGE, T/R RELAY, 10 dB PAD, LPF, PA LEADS, GATE BIAS SWITCH (continued)
USB HUB TUSB2046B, PORT TERMINATIONS, SPARE PORT
page 2 of 5 MeshSat field kit V2, CERN-OHL-S-2.0 PROTOTYPE, nothing built 2026-09-16
JST-PH 1x2 socket
TUSB2046BI four-port USB 2.0 full-..
6 MHz 3225
JST-PH 1x4 socket
USB AUDIO CODEC PCM2912A, HEADPHONE AMPLIFIER, MIC PREAMP, HEADSET LEADS
page 3 of 5 MeshSat field kit V2, CERN-OHL-S-2.0 PROTOTYPE, nothing built 2026-09-16
TI PCM2912A USB audio codec
decoupling of U6
TI TPA6132A2 headphone amplifier
TLV9062IDGK dual op amp
p1,5
USB AUDIO CODEC PCM2912A, HEADPHONE AMPLIFIER, MIC PREAMP, HEADSET LEADS | PTT AND EMCON LOGIC, PTT MIRROR, LEDS, EXPANDER 0x26 WITH LEVEL STAGES, TEST POINTS, FLAGS
USB AUDIO CODEC PCM2912A, HEADPHONE AMPLIFIER, MIC PREAMP, HEADSET LEADS (continued)
PTT AND EMCON LOGIC, PTT MIRROR, LEDS, EXPANDER 0x26 WITH LEVEL STAGES, TEST POINTS, FLAGS

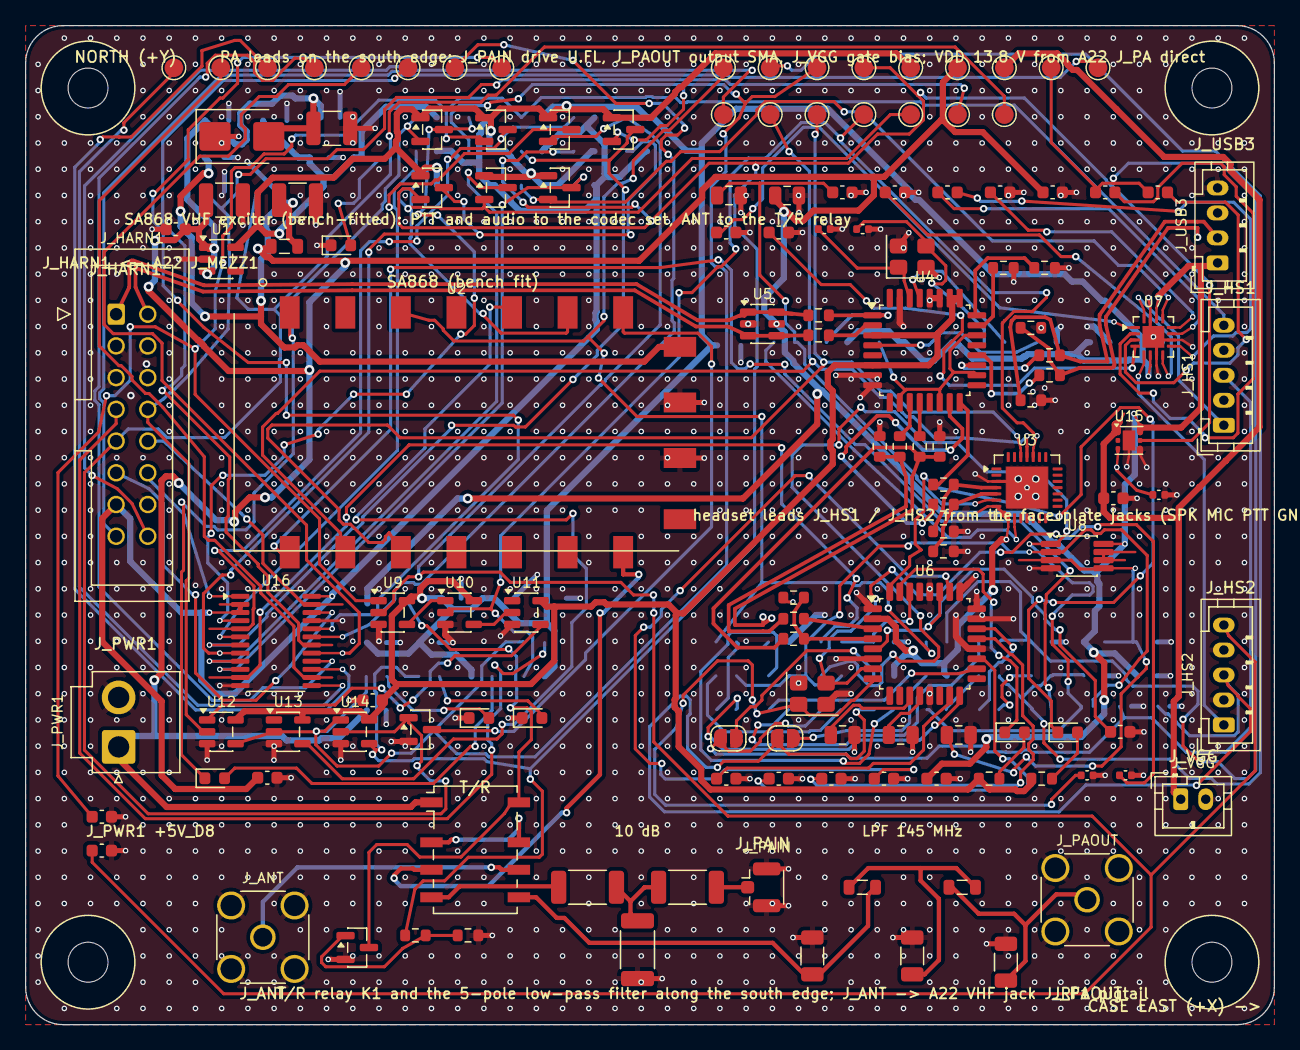
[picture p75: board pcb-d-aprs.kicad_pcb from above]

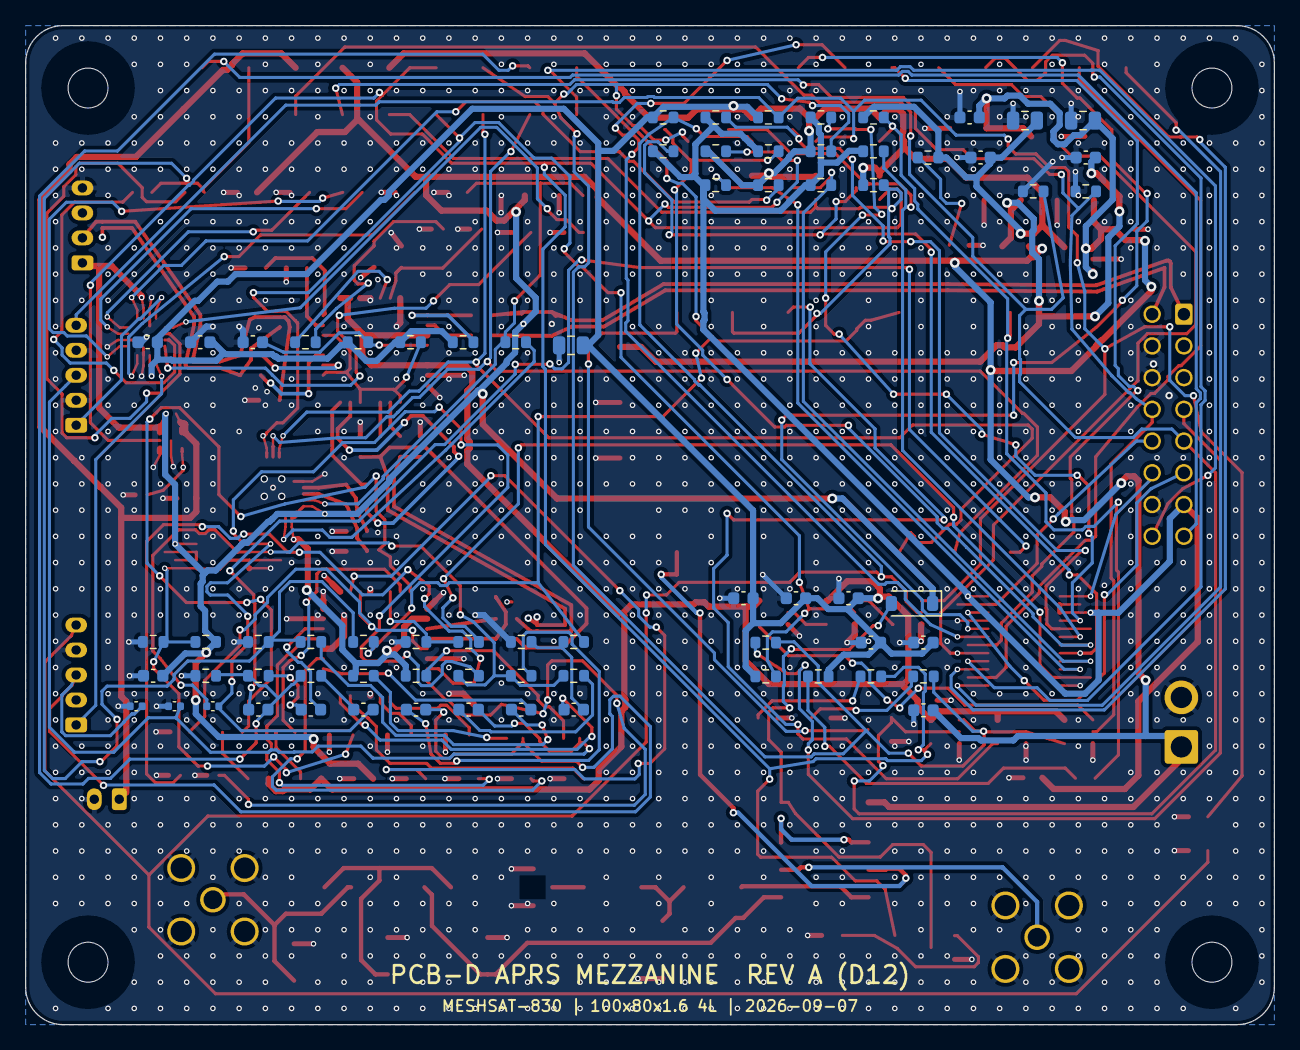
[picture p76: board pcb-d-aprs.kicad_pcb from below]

Board: 4 copper layers, 100.0 x 80.0 mm, 211 parts (71 on the bottom side), 133 nets.

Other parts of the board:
H1, H2, H3, H4: M3 standoff on A22 (5/95, +-35); MountingHole_3.2mm_M3

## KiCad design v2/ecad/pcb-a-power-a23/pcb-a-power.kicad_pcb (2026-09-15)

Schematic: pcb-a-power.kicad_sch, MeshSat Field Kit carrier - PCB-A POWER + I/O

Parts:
C1, C2: 47u 25V; C_1206_3216Metric
C3, C29, C30, C35, C36, C41, C42, C47, C48, C54, C120: 10u 25V 1210; C_1210_3225Metric
C4, C19: 1u; C_0603_1608Metric
C5, C26, C53, C57, C68, C75, C86, C98, C100, C102: 10n; C_0603_1608Metric
C6, C58, C69, C76, C87: 100p; C_0603_1608Metric
C7, C59, C70, C77, C88: 47n; C_0603_1608Metric
C8, C60, C71, C78, C89: 4.7u; C_0805_2012Metric
C9, C10, C16, C17, C61, C62, C72, C73, C79, C80, C90, C91: 100n 25V; C_0603_1608Metric
C11, C12, C13, C14, C15, C63, C64, C65, C66, C67, C74, C81, C82, C92, C108, C109, C110, C111, C116, C117, C118, C119: 10u 50V X7R 1210; C_1210_3225Metric
C18: 3.3u; C_0805_2012Metric
C20, C21, C22: 10u 35V 1210; C_1210_3225Metric
C23, C24, C25: 22u 25V 1210; C_1210_3225Metric
C27: 1n; C_0603_1608Metric
C28, C34, C40, C46, C52, C93, C95, C99, C101, C103, C104, C106, C107: 100n; C_0603_1608Metric
C31, C32, C33, C37, C38, C39, C43, C44, C45, C49, C50, C51, C55, C56: 22u 10V X7R 1210; C_1210_3225Metric
C83, C84, C85: 10u 100V X7R 1210; C_1210_3225Metric
C94: 220n; C_0603_1608Metric
C96, C97: 330p; C_0603_1608Metric
C112, C113, C114, C115: 3.3n; C_0603_1608Metric
D1: SMCJ18A (VBAT clamp); D_SMC; LCSC C374030
D2: SMCJ33A (VIN_RAW clamp behind E6's filter); D_SMC
D3: SMBJ5.0A; D_SMB
D4: SMBJ18A (VBUS clamp at the outlet); D_SMB
F1: 25 A mini blade (Keystone 3568 holder): pack node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; Fuseholder_Blade_Mini_Keystone_3568
J_5V_DEV: USB device rail to B16 (JST-VH): + -; JST_VH_B2P-VH_1x02_P3.96mm_Vertical; LCSC C274411
J_5V_S1: slot 1 5.1 V rail to B16 (JST-VH, 16 AWG): + -; JST_VH_B2P-VH_1x02_P3.96mm_Vertical; LCSC C274411
J_5V_S2: slot 2 5.1 V rail to B16 (JST-VH, 16 AWG): + -; JST_VH_B2P-VH_1x02_P3.96mm_Vertical; LCSC C274411
J_5V_S3: slot 3 5.1 V rail to B16 (JST-VH, 16 AWG): + -; JST_VH_B2P-VH_1x02_P3.96mm_Vertical; LCSC C274411
J_54V: 54 V to the PoE injector on B16 (JST-VH): + -; JST_VH_B2P-VH_1x02_P3.96mm_Vertical; LCSC C274411
J_AB1: A-B interconnect (IDC 2x13, top side) to B16's un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; IDC-Header_2x13_P2.54mm_Vertical_NarrowPad
J_AB2: A-B wall-port ribbon (IDC 2x5): the wall USB pair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; IDC-Header_2x05_P2.54mm_Vertical_NarrowPad
J_BM1, J_BM2, J_BM3, J_BM4, J_BM5, J_BM6, J_BM7, J_BM8, J_BM9, J_BM10, J_BM11: SMP-MAX slide-on receptacle R222M00720 (underside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; Radiall_SMPMAX_R222M00720
J_CN1, J_CN2, J_CN3, J_CN4: 9 A spring pin, pack return (Mill-Max 0858 class,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; Mill-Max_0858_power_pin
J_CP1, J_CP2, J_CP3, J_CP4: 9 A spring pin, CELL+ (Mill-Max 0858 class, dock 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; Mill-Max_0858_power_pin
J_DOCK: spring pins to the dock block (2x6, Preci-Dip 813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; PogoPins_2x6
J_HEAT: JST-XH 1x2 socket: the heater mat under the 2590 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; JST_XH_B2B-XH-A_1x02_P2.50mm_Vertical; LCSC C265283
J_HF: 12.0 V to the QMX HF unit in its lid tray (JST-VH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; JST_VH_B2P-VH_1x02_P3.96mm_Vertical; LCSC C274411
J_MAINSW: JST-XH 1x2 socket: the MAIN button lead from the 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; JST_XH_B2B-XH-A_1x02_P2.50mm_Vertical; LCSC C265283
J_MEZZ1: D8 mezzanine harness (IDC 2x8): its USB pair, the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; IDC-Header_2x08_P2.54mm_Vertical_NarrowPad
J_MEZZ_PWR1: D8 mezzanine 5 V (JST-VH): + -; JST_VH_B2P-VH_1x02_P3.96mm_Vertical; LCSC C274411
J_MON: monitor supply lead to the Xenarc (JST-VH): + -; JST_VH_B2P-VH_1x02_P3.96mm_Vertical; LCSC C274411
J_PA: 13.8 V to the PA module on the face plate (JST-VH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; JST_VH_B2P-VH_1x02_P3.96mm_Vertical; LCSC C274411
J_PRE1: pre-charge pin, longer, mates first (32.24 AX); Mill-Max_0858_power_pin
J_RF1, J_RF2, J_RF3, J_RF4, J_RF5, J_RF6, J_RF7, J_RF8, J_RF9, J_RF10, J_RF11: SMA jack, Amphenol 132134-11 vertical (pigtail to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; SMA_Amphenol_132134-11_Vertical; LCSC C3174425
J_USBC_OUT: wall USB-C outlet, power side (pigtail header): V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; PinHeader_1x05_P2.54mm_Vertical
J_USBW: JST-PH 1x4 socket: the wall USB-C data pair to B1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; JST_PH_B4B-PH-K_1x04_P2.00mm_Vertical; LCSC C131334
L1: 10uH XAL1010-103ME (Isat 14 A); L_Coilcraft_XAL1010-XXX
L2: 3.3uH XAL6030-332ME (Isat 12.2 A); L_Coilcraft_XAL6060-XXX
L3, L4, L5, L6: 4.7uH XAL6060-472ME (Isat 11 A); L_Coilcraft_XAL6060-XXX
L7: 4.7uH XAL4030-472ME; L_Coilcraft_XAL4030-XXX
L8: 6.8uH XAL1010-682ME (Isat 17 A); L_Coilcraft_XAL1010-XXX
L9, L11: 6.8uH XAL1010-682ME; L_Coilcraft_XAL1010-XXX
L10: 22uH XAL1010-223ME (Isat 9 A); L_Coilcraft_XAL1010-XXX
Q1: 2N7002: panel controller high = pull KILL low = p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; SOT-23
Q2, Q3, Q4, Q5, Q17, Q18, Q19, Q20: CSD19532Q5B 100 V N-FET (4.6 mOhm at VGS 6 V, Pow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; PowerPAK_SO-8_Single; LCSC C473333
Q6: 2N7002: CHG_INHIBIT high = ILIM_HIZ low = charger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; SOT-23
Q7, Q8, Q9, Q10, Q11, Q12, Q13, Q14, Q15, Q16, Q21, Q22, Q23, Q24, Q25, Q26: CSD18510Q5B 40 V N-FET; PowerPAK_SO-8_Single
Q27: CSD18510Q5B 40 V N-FET (VBUS switch); PowerPAK_SO-8_Single
R1: 10R 2W 2512; R_2512_6332Metric
R2, R3, R4, R5, R13, R21, R30, R34, R38, R42, R57, R73, R102, R103, R104, R111, R112, R113, R114, R116, R118, R123, R128, R143, R145: 100k; R_0603_1608Metric
R6: 240k 1%; R_0603_1608Metric
R7, R15, R29, R33, R37, R41, R49, R51, R59, R61, R67, R75, R125, R134: 10k 1%; R_0603_1608Metric
R8, R52, R62, R68, R78: 40.2k (300 kHz); R_0603_1608Metric
R9, R53, R63, R69, R79: 30k (slope); R_0603_1608Metric
R10, R22, R23, R25, R44, R54, R64, R70, R80, R91, R95, R99, R110, R117, R142: 10k; R_0603_1608Metric
R11, R65, R81, R138: 10mOhm 1% 2512 (ISNS); R_2512_6332Metric
R12, R56, R122, R127: 5mOhm 1% 2512 (CS); R_2512_6332Metric
R14, R58, R74, R124, R133: 62k 1%; R_0603_1608Metric
R16: 10mOhm 1% 2512 (RAC, input current sense); R_2512_6332Metric
R17: 5mOhm 1% 2512 (RSR, charge current sense); R_2512_6332Metric
R18: 10R; R_0603_1608Metric
R19: 16.5k 1%; R_0603_1608Metric
R20: 34.8k 1%; R_0603_1608Metric
R24: 10k (PSYS load); R_0603_1608Metric
R26: 60.4k 1% (CELL_BATPRESZ: 4S per Table, from VDDA); R_0603_1608Metric
R27: 40.2k 1%; R_0603_1608Metric
R28, R32, R36, R40: 53.6k 1%; R_0603_1608Metric
R31, R35, R39, R43: 5mOhm 1% 2512 (shunt); R_2512_6332Metric
R45, R46, R47, R115: 68k (RT: 500 kHz); R_0603_1608Metric
R48: 31.6k 1%; R_0603_1608Metric
R50: 162k 1%; R_0603_1608Metric
R55: 2mOhm 1% 2512 (ISNS); R_2512_6332Metric
R60: 140k 1%; R_0603_1608Metric
R66: 665k 1%; R_0603_1608Metric
R71: 20mOhm 1% 2512 (ISNS); R_2512_6332Metric
R72: 10mOhm 1% 2512 (CS); R_2512_6332Metric
R76: 105k 1%; R_0603_1608Metric
R77: 20k 1% (R_FBL); R_0603_1608Metric
R90: 750R 1% (ILM: 1.2 A); R_0603_1608Metric
R92, R96, R100: 100k 1%; R_0603_1608Metric
R93, R97, R101: 10k 1% (OVLO); R_0603_1608Metric
R94: 909R 1% (ILM: 1.0 A); R_0603_1608Metric
R98: 453R 1% (ILM: 2.0 A); R_0603_1608Metric
R119, R120, R121, R126, R135: 100k (MODE: CCM); R_0603_1608Metric
R129, R130, R131, R132: 22k; R_0603_1608Metric
R136: 21.0k 1% (R_FBL2: 9 V when CTL2 is low); R_0603_1608Metric
R137: 14.0k 1% (R_FBL1: 15 V when CTL1 is low too); R_0603_1608Metric
R139: 43R 1W 2512 (DSCG); R_2512_6332Metric
R140: 1M (GD to VPWR, 9.1.3); R_0603_1608Metric
R141: 698k; R_0603_1608Metric
TP3: EXP2_SP3; TestPoint_Pad_D1.5mm
TP4: EXP2_SP4; TestPoint_Pad_D1.5mm
TP5: EXP2_SP5; TestPoint_Pad_D1.5mm
TP6: EXP2_SP6; TestPoint_Pad_D1.5mm
TP7: EXP2_SP7; TestPoint_Pad_D1.5mm
TP8: EXP2_SP8; TestPoint_Pad_D1.5mm
TP9: VBAT; TestPoint_Pad_D1.5mm
TP10: GND; TestPoint_Pad_D1.5mm
TP11: +3V3; TestPoint_Pad_D1.5mm
TP12: VBUS20; TestPoint_Pad_D1.5mm
TP13: VIN_RAW; TestPoint_Pad_D1.5mm
TP14: CELL+; TestPoint_Pad_D1.5mm
TP15: EMCON_HW; TestPoint_Pad_D1.5mm
TP16: RAIL_EN; TestPoint_Pad_D1.5mm
TP17: SDA; TestPoint_Pad_D1.5mm
TP18: SCL; TestPoint_Pad_D1.5mm
TP19: IADPT; TestPoint_Pad_D1.5mm
TP20: IBAT; TestPoint_Pad_D1.5mm
TP21: DOCK_SPARE; TestPoint_Pad_D1.5mm
TP22: REGN; TestPoint_Pad_D1.5mm
TP23: EXP2_SPA; TestPoint_Pad_D1.5mm
TP24: EXP2_SPB; TestPoint_Pad_D1.5mm
TP25: EXP2_SPC; TestPoint_Pad_D1.5mm
TP26: EXP2_SPD; TestPoint_Pad_D1.5mm
TP27: AB_SPARE; TestPoint_Pad_D1.5mm
U1: LTC2954CTS8-1 push-button on/off controller; TSOT-23-8; LCSC C683782
U2: LM5176PWPR buck-boost controller, VBUS20 from VIN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; HTSSOP-28-1EP_4.4x9.7mm_P0.65mm_EP2.85x5.4mm; LCSC C442493
U3: BQ25731RSNR 1 to 5 cell buck-boost charger, 4S fr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; QFN-32-1EP_4x4mm_P0.4mm_EP2.65x2.65mm; LCSC C2871872
U4: AP64500SP-13 5 A buck, 5.1 V rail +5V_S1; SOIC-8-1EP_3.9x4.9mm_P1.27mm_EP2.29x3mm; LCSC C2070920
U5: AP64500SP-13 5 A buck, 5.1 V rail +5V_S2; SOIC-8-1EP_3.9x4.9mm_P1.27mm_EP2.29x3mm; LCSC C2070920
U6: AP64500SP-13 5 A buck, 5.1 V rail +5V_S3; SOIC-8-1EP_3.9x4.9mm_P1.27mm_EP2.29x3mm; LCSC C2070920
U7: AP64500SP-13 5 A buck, 5.1 V rail +5V_DEV; SOIC-8-1EP_3.9x4.9mm_P1.27mm_EP2.29x3mm; LCSC C2070920
U8: INA226 rail monitor +5V_S1; VSSOP-10_3x3mm_P0.5mm; LCSC C49851
U9: INA226 rail monitor +5V_S2; VSSOP-10_3x3mm_P0.5mm; LCSC C49851
U10: INA226 rail monitor +5V_S3; VSSOP-10_3x3mm_P0.5mm; LCSC C49851
U11: INA226 rail monitor +5V_DEV; VSSOP-10_3x3mm_P0.5mm; LCSC C49851
U12: TPS62933DRLR 3 A buck, 3.3 V logic; SOT-583-8; LCSC C3200405
U13: LM5176PWPR buck-boost controller, +13V8_PA from V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; HTSSOP-28-1EP_4.4x9.7mm_P0.65mm_EP2.85x5.4mm; LCSC C442493
U14: INA226 PA rail monitor (0x46); VSSOP-10_3x3mm_P0.5mm; LCSC C49851
U15: LM5176PWPR buck-boost controller, +12V_HF from VB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; HTSSOP-28-1EP_4.4x9.7mm_P0.65mm_EP2.85x5.4mm; LCSC C442493
U16: LM5176PWPR buck-boost controller, +54V_POE from V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; HTSSOP-28-1EP_4.4x9.7mm_P0.65mm_EP2.85x5.4mm; LCSC C442493
U17: INA226 PoE rail monitor (0x47); VSSOP-10_3x3mm_P0.5mm; LCSC C49851
U18: TPS25740ARGER USB-C PD source controller, 45 W ou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; QFN-24-1EP_4x4mm_P0.5mm_EP2.5x2.5mm; LCSC C544309
U19: LM5176PWPR buck-boost controller, PD_VPWR from VB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; HTSSOP-28-1EP_4.4x9.7mm_P0.65mm_EP2.85x5.4mm; LCSC C442493
U21: TPS259631DDAR eFuse VBAT -> VMON (750R 1% (ILM: 1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; SOIC-8-1EP_3.9x4.9mm_P1.27mm_EP2.29x3mm; LCSC C2155778
U22: TPS259631DDAR eFuse VBAT -> VHEAT (909R 1% (ILM: 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; SOIC-8-1EP_3.9x4.9mm_P1.27mm_EP2.29x3mm; LCSC C2155778
U23: TPS259631DDAR eFuse +5V_DEV -> +5V_D8 (453R 1% (I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; SOIC-8-1EP_3.9x4.9mm_P1.27mm_EP2.29x3mm; LCSC C2155778
U26: SN74LVC08APWR quad AND: EMCON gates for the PA ra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; TSSOP-14_4.4x5mm_P0.65mm; LCSC C465737
U27: PCA9555PW (0x21): enables and status; TSSOP-24_4.4x7.8mm_P0.65mm; LCSC C2864778
U28: PCA9555PW (0x24): power-good lines, spares; TSSOP-24_4.4x7.8mm_P0.65mm; LCSC C2864778
U29: USBLC6-2SC6; SOT-23-6; LCSC C7519
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

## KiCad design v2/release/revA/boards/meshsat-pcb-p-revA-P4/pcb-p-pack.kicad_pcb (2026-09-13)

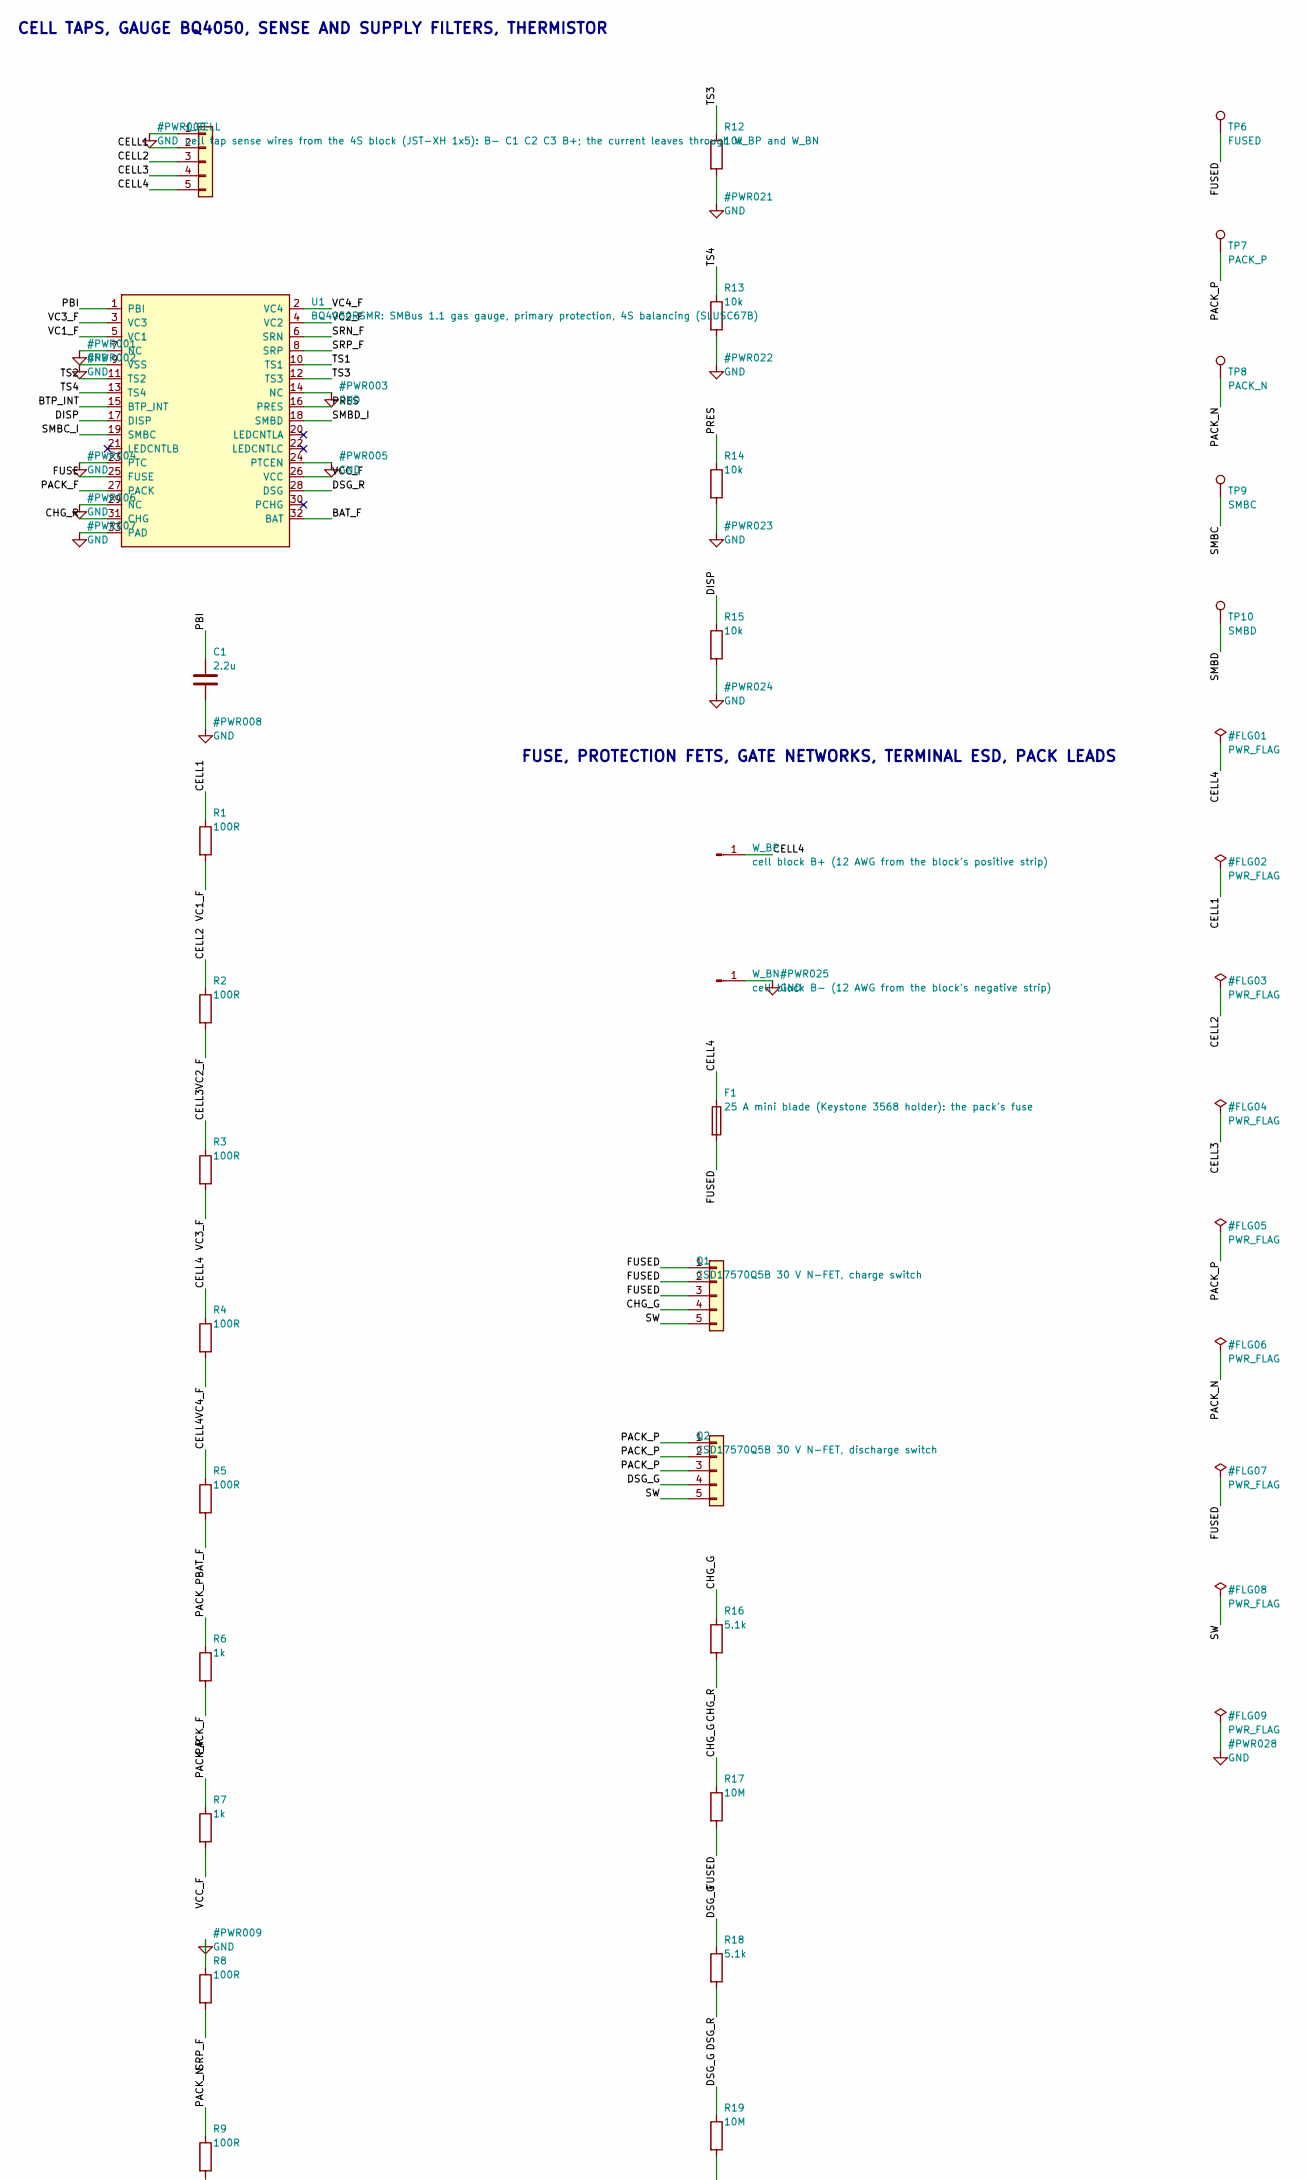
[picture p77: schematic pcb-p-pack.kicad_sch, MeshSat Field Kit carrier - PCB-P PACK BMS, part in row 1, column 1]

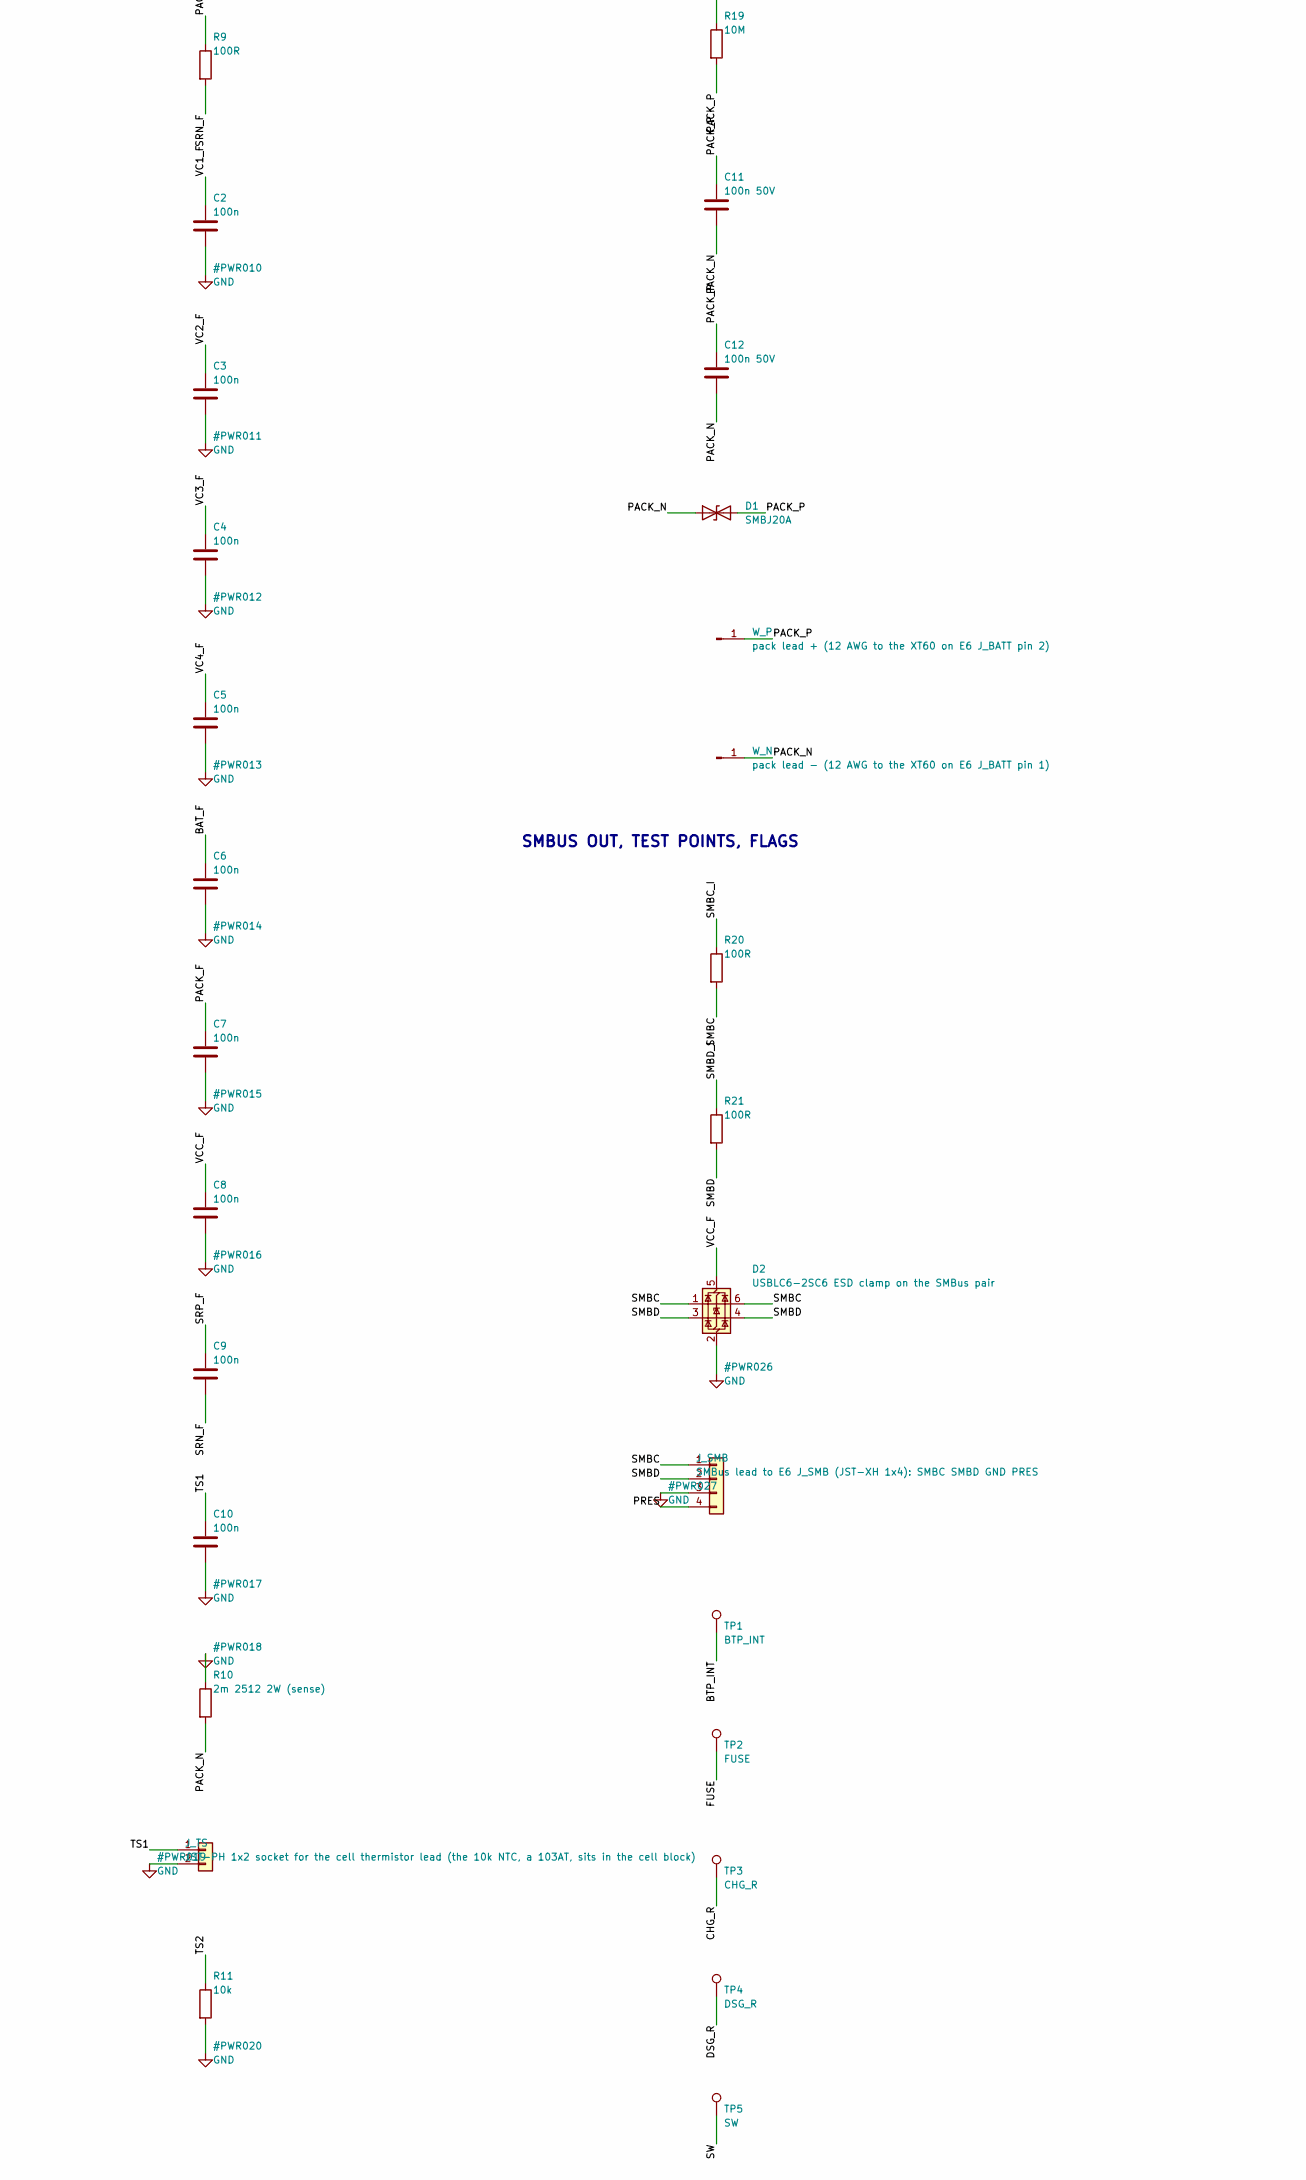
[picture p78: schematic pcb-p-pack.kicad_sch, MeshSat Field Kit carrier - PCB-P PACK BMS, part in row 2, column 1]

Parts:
C1: 2.2u; C_0805_2012Metric
C2, C3, C4, C5, C6, C7, C8, C9, C10: 100n; C_0603_1608Metric
C11: 100n 50V; C_0603_1608Metric
C12: 100n 50V; C_1206_3216Metric
D1: SMBJ20A; D_SMB
D2: USBLC6-2SC6 ESD clamp on the SMBus pair; SOT-23-6; LCSC C7519
F1: 25 A mini blade (Keystone 3568 holder): the pack'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; Fuseholder_Blade_Mini_Keystone_3568
J_CELL: cell tap sense wires from the 4S block (JST-XH 1x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; JST_XH_B5B-XH-A_1x05_P2.50mm_Vertical
J_SMB: SMBus lead to E6 J_SMB (JST-XH 1x4): SMBC SMBD GN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; JST_XH_B4B-XH-A_1x04_P2.50mm_Vertical
J_TS: JST-PH 1x2 socket for the cell thermistor lead (t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; JST_PH_B2B-PH-K_1x02_P2.00mm_Vertical; LCSC C5251182
Q1: CSD17570Q5B 30 V N-FET, charge switch; PowerPAK_SO-8_Single; LCSC C529279
Q2: CSD17570Q5B 30 V N-FET, discharge switch; PowerPAK_SO-8_Single; LCSC C529279
R1, R2, R3, R4, R5, R8, R9, R20, R21: 100R; R_0603_1608Metric
R6, R7: 1k; R_0603_1608Metric
R10: 2m 2512 2W (sense); R_2512_6332Metric
R11, R12, R13, R14, R15: 10k; R_0603_1608Metric
R16, R18: 5.1k; R_0603_1608Metric
R17, R19: 10M; R_0603_1608Metric
TP1: BTP_INT; TestPoint_Pad_D1.5mm
TP2: FUSE; TestPoint_Pad_D1.5mm
TP3: CHG_R; TestPoint_Pad_D1.5mm
TP4: DSG_R; TestPoint_Pad_D1.5mm
TP5: SW; TestPoint_Pad_D1.5mm
TP6: FUSED; TestPoint_Pad_D1.5mm
TP7: PACK_P; TestPoint_Pad_D1.5mm
TP8: PACK_N; TestPoint_Pad_D1.5mm
TP9: SMBC; TestPoint_Pad_D1.5mm
TP10: SMBD; TestPoint_Pad_D1.5mm
U1: BQ4050RSMR: SMBus 1.1 gas gauge, primary protecti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; QFN-32-1EP_5x5mm_P0.5mm_EP3.1x3.1mm; LCSC C157570
W_BN: cell block B- (12 AWG from the block's negative s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; SolderWire-2.5sqmm_1x01_D2.4mm_OD3.6mm
W_BP: cell block B+ (12 AWG from the block's positive s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; SolderWire-2.5sqmm_1x01_D2.4mm_OD3.6mm
W_N: pack lead - (12 AWG to the XT60 on E6 J_BATT pin 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; SolderWire-2.5sqmm_1x01_D2.4mm_OD3.6mm
W_P: pack lead + (12 AWG to the XT60 on E6 J_BATT pin 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; SolderWire-2.5sqmm_1x01_D2.4mm_OD3.6mm

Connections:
/BAT_F: C6.1, R5.2, U1.32 (BAT)
/BTP_INT: TP1.1, U1.15 (BTP_INT)
/CELL1: J_CELL.2, R1.1
/CELL2: J_CELL.3, R2.1
/CELL3: J_CELL.4, R3.1
/CELL4: F1.1, J_CELL.5, R4.1, R5.1, W_BP.1
/CHG_G: Q1.4, R16.1, R17.1
/CHG_R: R16.2, TP3.1, U1.31 (CHG)
/DISP: R15.1, U1.17 (DISP)
/DSG_G: Q2.4, R18.1, R19.1
/DSG_R: R18.2, TP4.1, U1.28 (DSG)
/FUSE: TP2.1, U1.25 (FUSE)
/FUSED: F1.2, Q1.1, Q1.2, Q1.3, R17.2, TP6.1
/PACK_F: C7.1, R6.2, U1.27 (PACK)
/PACK_N: C11.2, C12.2, D1.1 (A1), R9.1, R10.2, TP8.1, W_N.1
/PACK_P: C11.1, C12.1, D1.2 (A2), Q2.1, Q2.2, Q2.3, R6.1, R7.1, R19.2, TP7.1, W_P.1
/PBI: C1.1, U1.1 (PBI)
/PRES: J_SMB.4, R14.1, U1.16 (PRES)
/SMBC: D2.1 (I/O1), D2.6 (I/O1), J_SMB.1, R20.2, TP9.1
/SMBC_I: R20.1, U1.19 (SMBC)
/SMBD: D2.3 (I/O2), D2.4 (I/O2), J_SMB.2, R21.2, TP10.1
/SMBD_I: R21.1, U1.18 (SMBD)
/SRN_F: C9.2, R9.2, U1.6 (SRN)
/SRP_F: C9.1, R8.2, U1.8 (SRP)
/SW: Q1.5, Q2.5, TP5.1
/TS1: C10.1, J_TS.1, U1.10 (TS1)
/TS2: R11.1, U1.11 (TS2)
/TS3: R12.1, U1.12 (TS3)
/TS4: R13.1, U1.13 (TS4)
/VC1_F: C2.1, R1.2, U1.5 (VC1)
/VC2_F: C3.1, R2.2, U1.4 (VC2)
/VC3_F: C4.1, R3.2, U1.3 (VC3)
/VC4_F: C5.1, R4.2, U1.2 (VC4)
/VCC_F: C8.1, D2.5 (VBUS), R7.2, U1.26 (VCC)
GND: C1.2, C2.2, C3.2, C4.2, C5.2, C6.2, C7.2, C8.2, C10.2, D2.2 (GND), J_CELL.1, J_SMB.3, J_TS.2, R8.1, R10.1, R11.2, R12.2, R13.2, R14.2, R15.2, U1.7 (NC), U1.9 (VSS), U1.14 (NC), U1.23 (PTC), U1.24 (PTCEN), U1.29 (NC), U1.33 (PAD), W_BN.1

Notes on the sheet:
CELL TAPS, GAUGE BQ4050, SENSE AND SUPPLY FILTERS, THERMISTOR
FUSE, PROTECTION FETS, GATE NETWORKS, TERMINAL ESD, PACK LEADS
SMBUS OUT, TEST POINTS, FLAGS

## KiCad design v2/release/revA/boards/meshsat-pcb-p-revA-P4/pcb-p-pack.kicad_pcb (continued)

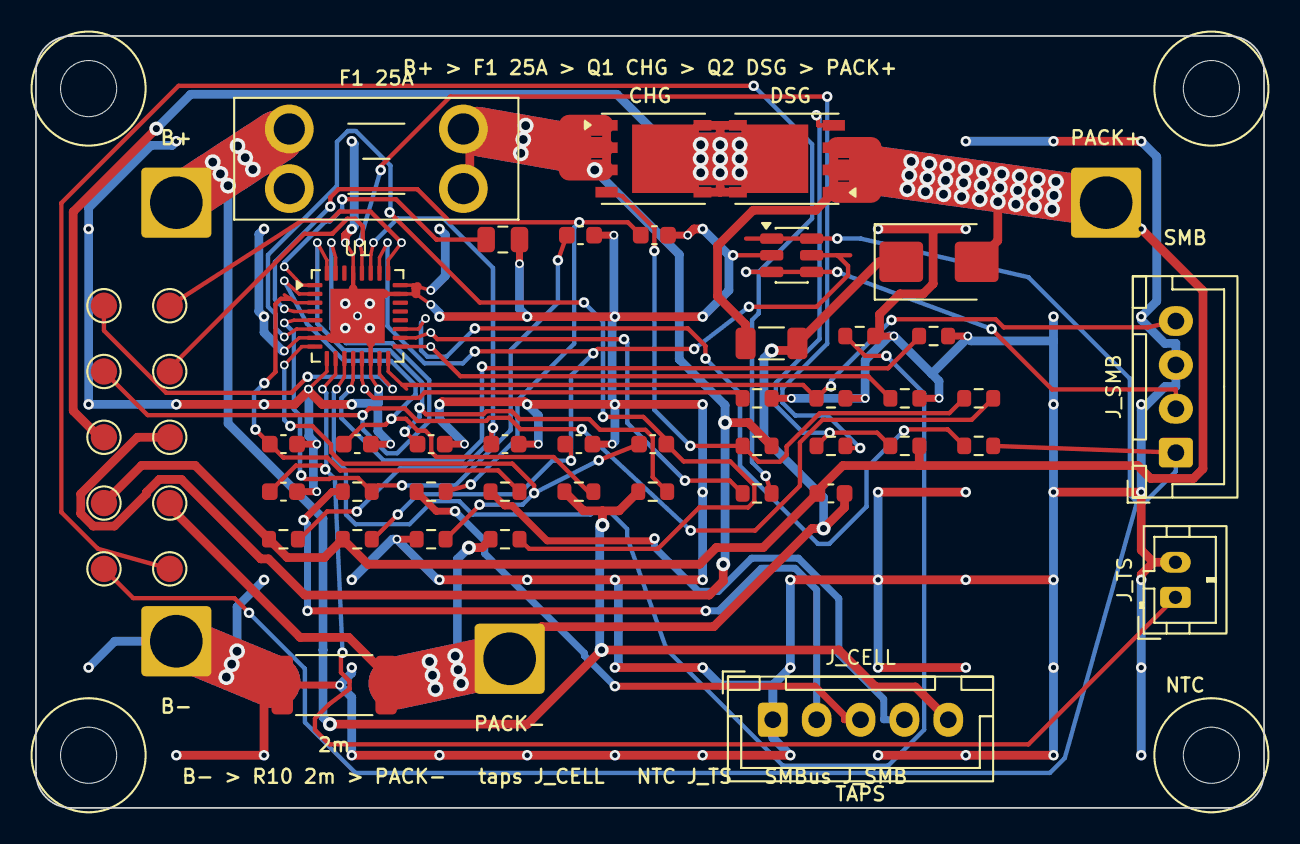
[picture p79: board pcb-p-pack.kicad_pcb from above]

Board: 2 copper layers, 70.0 x 44.0 mm, 60 parts (0 on the bottom side), 35 nets.

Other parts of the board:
H1, H2, H3, H4: M3 into the enclosure boss; MountingHole_3.2mm_M3

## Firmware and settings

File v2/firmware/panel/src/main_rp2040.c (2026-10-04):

/*
 * main_rp2040.c: the panel controller's main loop on the RP2040 (pico-sdk). NOT BUILT HERE (no arm toolchain on this
 * host); prototype firmware for an unbuilt board.
 *
 * Order (FW-C01, FW-C02): PI_KILL low and PI_SHDN_REQ released first; ZEROIZE_SW and the SLOT_EN pads read as inputs;
 * the core decides each SLOT_EN's first level (all low with the toggle closed or a wipe pending); the watchdog; then
 * the 1 ms loop, in which the core runs the rest of the boot order (the wipe table, the expanders, the charger (owed),
 * HOT-R1, the slots one at a time).
 *
 * Not here, and owed (README.md section 4): the USB device and the bridge protocol (MESHSAT-837, wire format not
 * defined), the e-paper's command layer, the charger's registers (FW-A rows), the secure element's command layer
 * (CryptoAuthLib, not vendored), the VEML7700 and TMP117 reads.
 */
#include <stdbool.h>

#include "hal.h"
#include "panel.h"

void hal_init_rest(void);

static panel_t P;

/* FW-K04: after a failed transfer, a held SDA is released by nine SCL pulses and a STOP, and the event is logged */
static void bb_scl(void *c, bool l) { (void)c; hal_i2c_bitbang_scl(l); }
static bool bb_sda(void *c) { (void)c; return hal_i2c_bitbang_sda_read(); }
static void bb_stop(void *c) { (void)c; hal_i2c_bitbang_stop(); }
static void bb_delay(void *c, unsigned us) { (void)c; hal_delay_us(us); }
static const panel_bitbang_t BB = { 0, bb_scl, bb_sda, bb_stop, bb_delay };

static int recover_if_held(int r)
{
    if (r == 0)
        return 0;
    hal_i2c_bitbang_begin();
    if (!hal_i2c_bitbang_sda_read()) {
        int pulses = panel_bus_recover(&BB);
        panel_ev_report(&P, EV_I2C_RECOVERED, (uint8_t)(pulses < 0 ? 0xFF : pulses), hal_now_ms());
    }
    hal_i2c_bitbang_end();
    return r;
}

static int bus_write(void *ctx, uint8_t addr, const uint8_t *buf, unsigned len)
{
    (void)ctx;
    return recover_if_held(hal_i2c_write(addr, buf, len, hal_now_ms() + HAL_I2C_OP_TIMEOUT_MS));
}

static int bus_read(void *ctx, uint8_t addr, uint8_t reg, uint8_t *buf, unsigned len)
{
    (void)ctx;
    ms_t d = hal_now_ms() + HAL_I2C_OP_TIMEOUT_MS;
    if (hal_i2c_write(addr, &reg, 1, d) != 0)
        return recover_if_held(-1);
    return recover_if_held(hal_i2c_read(addr, buf, len, d));
}

static ms_t z_now(void *ctx) { (void)ctx; return hal_now_ms(); }

/* The secure element's two GenKey modes go through CryptoAuthLib (atcab_genkey, atcab_get_pubkey) with the panel's
 * six-function HAL bounded as ZEROIZE.md 3.4 (a) and (b) set out. The library is not vendored in this tree: OWED. Until
 * it is, every SE call fails, so the boot table takes "the SE does not answer" (normal boot without the SE, MASTER WARN)
 * and a ZEROIZE commit ends INCOMPLETE with the slots held off: fail secure. */
static int se_create(void *ctx, uint8_t slot, uint8_t pub[64], ms_t deadline)
{
    (void)ctx; (void)slot; (void)pub; (void)deadline;
    return -1;
}
static int se_public(void *ctx, uint8_t slot, uint8_t pub[64], ms_t deadline)
{
    (void)ctx; (void)slot; (void)pub; (void)deadline;
    return -1;
}
static bool se_recorded(void *ctx, uint8_t slot, uint8_t pub[64])
{
    (void)ctx; (void)slot; (void)pub;
    return false;                            /* P_A0 and P_B0 are written at enrolment (ZEROIZE.md 3.3): owed */
}
static void arm_cut(void *ctx, ms_t at) { (void)ctx; hal_arm_slot_cut_alarm(at); }
static void tell_modules(void *ctx) { (void)ctx; /* over the bridge protocol: owed (F-02) */ }
static void feed(void *ctx) { (void)ctx; hal_watchdog_feed(); }
static int fl_read(void *ctx, uint32_t off, uint8_t *buf, unsigned len) { (void)ctx; return hal_journal_read(off, buf, len); }
static int fl_prog(void *ctx, uint32_t off, const uint8_t *buf, unsigned len) { (void)ctx; return hal_journal_program(off, buf, len); }
static int fl_erase(void *ctx) { (void)ctx; return hal_journal_erase(); }
static void epd_send(void *ctx, uint8_t page, bool full) { (void)ctx; (void)page; (void)full; /* owed */ }
static int ss_read(void *ctx, uint32_t off, uint8_t *buf, unsigned len) { (void)ctx; return hal_slotstore_read(off, buf, len); }
static int ss_prog(void *ctx, uint32_t off, const uint8_t *buf, unsigned len) { (void)ctx; return hal_slotstore_program(off, buf, len); }
static int ss_erase(void *ctx) { (void)ctx; return hal_slotstore_erase(); }

static const panel_ops_t OPS = {
    .bus = { 0, bus_write, bus_read },
    .zer = { 0, z_now, se_create, se_public, se_recorded, arm_cut, tell_modules, feed, fl_read, fl_prog, fl_erase,
             8192u },
    .epd = { 0, epd_send },
    .slots = { 0, ss_read, ss_prog, ss_erase, 4096u },
};

int main(void)
{
    hal_init_pins_first();                                   /* FW-C01 steps 1 and 2 */
    bool zer_closed = !hal_gpio_get(HAL_GPIO_ZEROIZE_SW);    /* step 3: the level, at the first instruction */
    bool held[3], drive[3];
    hal_slot_en_read(held);                                  /* FW-C02 */
    panel_init(&P, &OPS, hal_now_ms(), zer_closed, held, hal_reset_was_power_on(), drive);   /* FW-C05 (F-15) */
    hal_slot_en_drive_initial(drive);
    panel_ev_report(&P, EV_BOOT, (uint8_t)hal_reset_reason(), hal_now_ms());   /* FW-C02: the boot reason logged */
    hal_init_rest();
    hal_watchdog_start(PANEL_WATCHDOG_MS);

    panel_in_t in = { 0 };
    panel_out_t out;
    in.br.display_slot = -1;
    in.br.soc_pct = -1;
    ms_t last = hal_now_ms();
    for (;;) {
        ms_t now = hal_now_ms();
        if (now == last) {
            continue;
        }
        last = now;
        in.test_sw = hal_gpio_get(HAL_GPIO_TEST_SW);
        in.sos_sw = hal_gpio_get(HAL_GPIO_SOS_SW);
        in.zeroize_sw = hal_gpio_get(HAL_GPIO_ZEROIZE_SW);
        in.emcon_rd = hal_gpio_get(HAL_GPIO_EMCON_RD_R);
        in.tr_aprs = hal_gpio_get(HAL_GPIO_TR_APRS);
        in.exp_int = hal_gpio_get(HAL_GPIO_EXP_INT);
        in.hb[0] = hal_gpio_get(HAL_GPIO_HB1);
        in.hb[1] = hal_gpio_get(HAL_GPIO_HB2);
        in.hb[2] = hal_gpio_get(HAL_GPIO_HB3);
        in.pi_shdn_req = hal_gpio_get(HAL_GPIO_PI_SHDN_REQ);
        in.pi_button = false;                                /* HAL_PI_BUTTON_WIRED 0: finding F-01 */
        in.epd_busy = hal_gpio_get(HAL_GPIO_EPD_BUSY);
        in.rail_mv = hal_rail_sense_mv();

        panel_tick(&P, now, &in, &out);

        hal_gpio_put(HAL_GPIO_PI_KILL, out.pi_kill);
        hal_pi_shdn_req_assert(out.pi_shdn_assert);
        hal_gpio_put(HAL_GPIO_SLOT_EN1, out.slot_en[0]);
        hal_gpio_put(HAL_GPIO_SLOT_EN2, out.slot_en[1]);
        hal_gpio_put(HAL_GPIO_SLOT_EN3, out.slot_en[2]);
        hal_gpio_put(HAL_GPIO_HDMI_SEL1, out.hdmi_sel1);
        hal_gpio_put(HAL_GPIO_HDMI_SEL2, out.hdmi_sel2);
        hal_gpio_put(HAL_GPIO_SHORE_INHIBIT, out.shore_inhibit);
        hal_gpio_put(HAL_GPIO_EPD_PWR_n, !out.epd_power);
        hal_gpio_put(HAL_GPIO_LED_STAT, out.led_stat);
        hal_pwm_set_permille(HAL_GPIO_PANEL_PWM, out.pwm_permille);
        hal_pwm_set_permille(HAL_GPIO_PWM1, out.sounder ? 1000u : 0u);
        hal_watchdog_feed();
    }
}

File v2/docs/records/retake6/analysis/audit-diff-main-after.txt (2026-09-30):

retake6: the audit of main 6ec37197 (from evidence-main-6ec37197.tar) against the audit in the worktree after the re-take
before: 339 rows; classes {'AWAITING_REVALIDATION': 215, 'CURRENT_CANDIDATE': 62, 'DESK_REVIEW': 21, 'NO_EVIDENCE': 22, 'VALID_HISTORICAL': 19}; results {'FAIL': 44, 'INCONCLUSIVE': 88, 'NOT_APPLICABLE': 1, 'PASS': 206}; CURRENT_CANDIDATE 62 of which PASS 57
after: 339 rows; classes {'AWAITING_REVALIDATION': 213, 'CURRENT_CANDIDATE': 83, 'DESK_REVIEW': 21, 'NO_EVIDENCE': 22}; results {'FAIL': 40, 'INCONCLUSIVE': 89, 'NOT_APPLICABLE': 1, 'PASS': 209}; CURRENT_CANDIDATE 83 of which PASS 71

ROWS WHOSE RESULT CHANGED
  A  RF-002   SCHEM FAIL         CURRENT_CANDIDATE (BOUND)  ->  INCONCLUSIVE CURRENT_CANDIDATE (BOUND)
       before: inhibit_chain_a FAIL: {'fail': 1, 'pass': 6, 'undecided': 2, 'unjudged': 0}
       after:  inhibit_chain_a INCONCLUSIVE: RF-002 on this board: where the transmit inhibit line runs, it is present, reaches the gate it keys, has the panel toggle as its only source, is buffered and no
  B  RF-002   SCHEM FAIL         CURRENT_CANDIDATE (BOUND)  ->  INCONCLUSIVE CURRENT_CANDIDATE (BOUND)
       before: inhibit_chain_b FAIL: {'fail': 11, 'pass': 6, 'undecided': 3, 'unjudged': 0}
       after:  inhibit_chain_b INCONCLUSIVE: RF-002 on this board: where the transmit inhibit line runs, it is present, reaches the gate it keys, has the panel toggle as its only source, is buffered and no
  C  PWR-001  SCHEM FAIL         VALID_HISTORICAL (RATIONALE)  ->  PASS         CURRENT_CANDIDATE (BOUND)
       before: intent_rails FAIL: {'census_nets': 153, 'checks': 7, 'declared_nodes': 1, 'declared_not_in_netlist': 0, 'declared_rails': 2, 'fail': 5, 'he
       after:  intent_rails PASS of 6
  C  RF-002   SCHEM FAIL         CURRENT_CANDIDATE (BOUND)  ->  PASS         CURRENT_CANDIDATE (BOUND)
       before: inhibit_chain_c FAIL: {'fail': 1, 'pass': 5, 'undecided': 0, 'unjudged': 0}
       after:  inhibit_chain_c PASS of 6
  D  PWR-001  SCHEM INCONCLUSIVE VALID_HISTORICAL (RATIONALE)  ->  PASS         CURRENT_CANDIDATE (BOUND)
       before: intent_rails INCONCLUSIVE: PWR-001 on the committed netlist and the intent file beside it: every power net is a declared rail, and every declared rail is a net of the netlist whose source
       after:  intent_rails PASS of 7
  D  RF-002   SCHEM FAIL         CURRENT_CANDIDATE (BOUND)  ->  INCONCLUSIVE CURRENT_CANDIDATE (BOUND)
       before: inhibit_chain_d FAIL: {'fail': 2, 'pass': 6, 'undecided': 0, 'unjudged': 0}
       after:  inhibit_chain_d INCONCLUSIVE: RF-002 on this board: where the transmit inhibit line runs, it is present, reaches the gate it keys, has the panel toggle as its only source, is buffered and no
  E  PWR-001  SCHEM INCONCLUSIVE VALID_HISTORICAL (RATIONALE)  ->  PASS         CURRENT_CANDIDATE (BOUND)
       before: intent_rails INCONCLUSIVE: PWR-001 on the committed netlist and the intent file beside it: every power net is a declared rail, and every declared rail is a net of the netlist whose source
       after:  intent_rails PASS of 16
  P  PWR-001  SCHEM FAIL         VALID_HISTORICAL (RATIONALE)  ->  PASS         CURRENT_CANDIDATE (BOUND)
       before: intent_rails FAIL: {'census_nets': 55, 'checks': 11, 'declared_nodes': 0, 'declared_not_in_netlist': 0, 'declared_rails': 5, 'fail': 6, 'he
       after:  intent_rails PASS of 11
  E5 SCH-003  ROUTE PASS         AWAITING_REVALIDATION (TOOL_CHANGED)  ->  FAIL         CURRENT_CANDIDATE (BOUND)
       before: check_contracts_e5 PASS of 33
       after:  check_contracts_e5 FAIL: {'fail': 10, 'pass': 28}
  E5 INT-001  SCHEM PASS         AWAITING_REVALIDATION (UNBOUND)  ->  FAIL         CURRENT_CANDIDATE (BOUND)
       before: interfaces_e5 PASS of 0
       after:  check_contracts_e5 FAIL: {'fail': 10, 'pass': 28}
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

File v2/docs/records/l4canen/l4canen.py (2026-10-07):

#!/usr/bin/env python3
"""l4canen.py: record l4canen, round 9 of record l9t5's task T10 (Layer 4 task L4A-54's correction on W139's quorum analysis, row (b)
of the AI-scope register; W143, MESHSAT-1357, 7 October 2026). PROTOTYPE DESIGN: nothing in this kit has been built, bought, powered
or measured; no figure printed here is a measurement.

It prints, deterministically and without touching the tree:
  1. the inputs, each pinned by sha256 (the makers' texts as the records' helper returns them);
  2. why: W139's finding W139-F2 (a supervisor latched off by W138's TPS2553-1 has nothing driving its EN) and the node W138 named;
  3. the composition on board B in L4-E9's change-list order with W137's canmb and W138's regstage in BOTH orders, with and without
     record l9t5's apply_gen_sch_b_canen.py after them: every step, the netlists equal in both orders, CON-004, canmb read by pin on
     the limiter's state, the limiter and regulator rows;
  4. the EN route read by pin, the mutations that must FAIL (an EN route a single peer can hold, among them) and the draft's refusals;
  5. the pin plan recounted (CON-017's convention) and read against DS12110 Table 9;
  6. the levels on the makers' printed rows (MODEL from PRINTED), the dark and faulty cases;
  7. the timing: the restart decision, the delay, the restart, the latched supervisor's RECOVERY INTERVAL, the rate and its energy;
  8. the route's own faults with their detection, and the route's in-service test riding on the restated self-test;
  9. FW-B21's stop at the loss count read against the corrected drafts, and the contract draft's text (DAR = 1 with ES0392's
     workaround quoted with its page, the restated self-test, the restart rule), composed on a scratch copy of the page;
 10. the SESSION decisions, the findings, what closes once independently checked;
 11. the predicates test_l4canen.py holds.
Run from the repository root:  python3 v2/docs/records/l4canen/l4canen.py  (about 20 s; it composes board B in temporary directories,
never the tree). Output: l4canen.out, regenerated with _bin/regen_out.py. Labels: PRINTED (a maker's limit), TYPICAL, DRAFTED (a
contract row or a drafted figure, not applied), MODEL, ASSUMPTION, SESSION."""
import ast
import hashlib
import importlib.util
import math
import os
import re
import shutil
import subprocess
import sys
import tempfile
import textwrap

HERE = os.path.dirname(os.path.abspath(__file__))
ROOT = os.path.dirname(os.path.dirname(os.path.dirname(os.path.dirname(HERE))))
sys.dont_write_bytecode = True
L9 = os.path.join(ROOT, "v2", "docs", "records", "l9t5")
sys.path.insert(0, L9)
import l9t5_canmb as M  # noqa: E402  (canmb's checks, CON-017's count and DS12110's Table 9 reader; its figures() is NOT called here)
D, CHK = M.D, M.CHK

# W34's convention (Q-41 item 1): every maker's text this record reads, each with its options; the held-back sheets' texts are held back
# with them (fetch_held_back.py beside this file). Re-take after a sheet changes: python3 v2/docs/records/_lib/retake_pdf_text.py
# v2/docs/records/l4canen
PDFTEXT = {
    "v2/vendor/power/aos-ao3400a-n-mosfet.pdf": [["-layout"]],
    "v2/vendor/st/st-es0392-rev15.pdf": [["-layout", "-f", "48", "-l", "48"]],
    "v2/vendor/st/st-rm0433-rev8.pdf": [["-layout", "-f", "533", "-l", "533"]],
    "v2/vendor/st/st-stm32h743xi-datasheet.pdf": [["-layout"]],
    "v2/vendor/ti/held/ti-tps2553-slvs841f.pdf": [["-layout"]],
    "v2/vendor/ti/held/ti-tps737-sbvs067w.pdf": [["-layout"]],
    "v2/vendor/ti/ti-sn74lvc1g08.pdf": [["-layout"]],
}
_PTS = importlib.util.spec_from_file_location("records_pdftext", os.path.join(ROOT, "v2", "docs", "records", "_lib", "pdftext.py"))
PDFT = importlib.util.module_from_spec(_PTS)
_PTS.loader.exec_module(PDFT)
REC = "v2/docs/records/l4canen"
SHEETS = {"fet": "v2/vendor/power/aos-ao3400a-n-mosfet.pdf", "es": "v2/vendor/st/st-es0392-rev15.pdf",
          "rm": "v2/vendor/st/st-rm0433-rev8.pdf", "h743": "v2/vendor/st/st-stm32h743xi-datasheet.pdf",
          "lim": "v2/vendor/ti/held/ti-tps2553-slvs841f.pdf", "ldo": "v2/vendor/ti/held/ti-tps737-sbvs067w.pdf",
          "g08": "v2/vendor/ti/ti-sn74lvc1g08.pdf"}
L9R = "v2/docs/records/l9t5"
DOCS = {"canen": L9R + "/apply_gen_sch_b_canen.py", "canmb": L9R + "/apply_gen_sch_b_canmb.py",
        "regstage": REC + "/inputs/l4reg-apply_gen_sch_b_regstage-469594bb.py", "sources": REC + "/inputs/SOURCES.txt",
        "guard": L9R + "/apply_gen_sch_b_iocguard.py", "iocset": L9R + "/apply_gen_sch_a_iocset.py", "iocpre": L9R + "/apply_gen_sch_b_iocpre.py",
        "canmb_py": L9R + "/l9t5_canmb.py", "canmb_out": L9R + "/l9t5_canmb.out", "canq_py": L9R + "/l9t5_canq.py",
        "canq_out": L9R + "/l9t5_canq.out", "canq_page": L9R + "/T10-CANQ.md", "contract": "v2/docs/HW-FW-CONTRACT.md",
        "contract_t10": L9R + "/apply_hw_fw_contract_t10.py", "contract_canq": L9R + "/apply_hw_fw_contract_canq.py",
        # W167 (W163-N4's class): l4reg_out is the tree's l4reg_compare.out (W159's envelope); it was L9R + "/inputs/l4reg-l4reg_compare-9fbda7a6.out"
        "l4reg_out": "v2/docs/records/l4reg/l4reg_compare.out", "drafts": L9R + "/l9t5_drafts.py",
        "gen_b": "v2/ecad/tools/gen_sch_b.py", "gennet": "v2/docs/records/l8p/gen_netlist.py", "trace": "v2/docs/REQUIREMENTS-TRACE.md"}
EN = chr(0x2013)       # the sheets' minus sign, written by its code point (no long dash in this file)
MU = "[%s%s]" % (chr(0xB5), chr(0x3BC))
TAGS = "ABC"
# DRAFTED by this round (the restart rule, apply_hw_fw_contract_canq.py) and SESSION (W143-D5): each printed with its reason in section 7
T_DEC = 2.0            # s: no edge on either of the target's TXDs and no state frame of it on either fabric for this long, at a peer
T_HOLD = 2.0           # s: a peer's restart vote is held this long, then released
T_RATE = 10.0          # s: at most one restart vote per target in this time (W139's route)
EN_LOW_MIN = 0.5       # s: the least time the route must hold the limiter's EN low (two orders over its printed turn-off time)
PULSE = (68e-3, 72e-3)     # s, a test pulse in the asserting peer's window (P1, P2 and V on the restart route)
READ = (66e-3, 74e-3)      # s, the target reads its restart gate's output over this span of its own window
# ASSUMPTION (a Layer 10 and Layer 6 part-selection bound, finding W143-F6): the RC's 4.7 uF keeps at least this much at 3.3 V over
# -20 to 85 C (21 % of nominal); its +10 % tolerance is the X7R class's, no part number being chosen yet
C_EFF_MIN, C_TOL = 1.0e-6, 0.10
C_RB_PF = 46.0         # ASSUMPTION, a Layer 10 bound: the read-back line, the reader's CIO included (as canmb's observation lines)
VGS_ON = 2.5           # V: the AO3400A's RDS(on) row is printed at this gate drive


def refuse(msg):
    sys.stderr.write("l4canen: REFUSED: %s\n" % msg)
    sys.exit(2)
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

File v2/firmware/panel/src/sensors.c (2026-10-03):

/*
 * sensors.c: the two kit-bus sensors the panel controller reads itself. Pure logic over the injected bus.
 *
 *  - Board B's TMP117 at 0x49 (FW-C13 and FW-C14's fallback with HOT-R1 held high). TI SNOSD82D (September 2022),
 *    held as v2/vendor/ti/ti-tmp117-temperature.pdf: the temperature register 00h is 16-bit two's complement at
 *    7.8125 m°C (section 7.6.2), reads 8000h (-256 °C) until the first conversion; the configuration register 01h
 *    resets to 0220h (continuous, 1 s cycle, 8 averages) and its bit 13 Data_Ready is set at the end of a conversion and
 *    cleared by a read of either register (Table 7-6). Registers are read MSB first. So a reading counts once per
 *    conversion: "two readings in a row" are two conversions, never one conversion read twice.
 *  - Board C's VEML7700 at 0x10 (P s.8: the reading reported to the bridge). Vishay 84286 Rev. 1.8 (28 November 2024),
 *    held as v2/vendor/vishay/veml7700-datasheet.pdf: ALS_CONF_0 (command 00h) powers up shut down (ALS_SD = 1);
 *    the firmware writes gain x1/8 (bits 12:11 = 10b) and 100 ms (bits 9:6 = 0000b), 1000h; ALS (04h) is 16 bit, LSB
 *    first. The lux per count at that setting is INFERRED by scaling the sheet's only printed figure, 0.0042 lx per step
 *    at gain x2 and 800 ms (lux = counts / (gain x responsivity), its Table 1 note): x16 for the gain, x8 for the
 *    time, 0.5376 lx per count; Vishay's application note, which the sheet refers to for the table, is not held.
 */
#include "panel.h"

#define TMP117_REG_TEMP 0x00
#define TMP117_REG_CONF 0x01
#define TMP117_DATA_READY (1u << 13)
#define TMP117_RESET_VALUE 0x8000u
#define VEML_ALS_CONF 0x00
#define VEML_ALS 0x04
#define VEML_CONF_GAIN_1_8_IT_100MS 0x1000u

int panel_tmp117_poll(panel_t *p, ms_t now)
{
    uint8_t b[2];
    p->tmp117_polled_at = now;
    if (p->ops->bus.i2c_read(p->ops->bus.ctx, HAL_I2C_TMP117, TMP117_REG_CONF, b, 2) != 0)
        goto fail;
    if (!(((unsigned)b[0] << 8 | b[1]) & TMP117_DATA_READY))
        return 0;                                            /* no new conversion since the last read */
    if (p->ops->bus.i2c_read(p->ops->bus.ctx, HAL_I2C_TMP117, TMP117_REG_TEMP, b, 2) != 0)
        goto fail;
    uint16_t raw = (uint16_t)((unsigned)b[0] << 8 | b[1]);
    if (raw == TMP117_RESET_VALUE)
        return 0;                                            /* before the first conversion */
    p->tmp117.valid = true;
    p->tmp117.mc = ((int32_t)(int16_t)raw * 125) / 16;        /* 7.8125 m°C a step */
    p->tmp117.seq++;
    p->tmp117_ok_at = now;
    return 0;
fail:
    if ((int32_t)(now - p->tmp117_ok_at) > 3000)
        p->tmp117.valid = false;                             /* no reading for 3 s: none */
    return -1;
}

int panel_veml_init(panel_t *p)
{
    uint8_t w[3] = { VEML_ALS_CONF, (uint8_t)(VEML_CONF_GAIN_1_8_IT_100MS & 0xFFu), (uint8_t)(VEML_CONF_GAIN_1_8_IT_100MS >> 8) };
    p->veml_ready = p->ops->bus.i2c_write(p->ops->bus.ctx, HAL_I2C_VEML7700, w, 3) == 0;
    return p->veml_ready ? 0 : -1;
}

int panel_veml_poll(panel_t *p, ms_t now)
{
    uint8_t b[2];
    p->veml_polled_at = now;
    if (!p->veml_ready && panel_veml_init(p) != 0)
        return -1;
    if (p->ops->bus.i2c_read(p->ops->bus.ctx, HAL_I2C_VEML7700, VEML_ALS, b, 2) != 0) {
        p->light_valid = false;
        p->veml_ready = false;                               /* re-written at the next poll (a power cycle shuts it down) */
        return -1;
    }
    p->light_counts = (uint16_t)(b[0] | (unsigned)b[1] << 8);
    p->light_mlux = (uint32_t)p->light_counts * 5376u / 10u; /* 0.5376 lx a count, INFERRED (header) */
    p->light_valid = true;
    return 0;
}

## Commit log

2026-09-28 chore(evidence): set 7's second re-take on the KiCad box at 05af085c after the tool fixes (the edge-rate readings re-taken with their note reworded; every schematic-phase reading current) [MESHSAT-13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
2026-09-28 docs(records): set 7's box logs filed (the second re-take's driver and writer logs, the suite at 7f6de345: 2171 passed, 0 failed, 3 skipped by host properties, and the two box helpers) [MESHSAT-1357]
2026-09-28 fix(records): stream energy: the unserved load is counted in every stopped hour (it was counted only at the stopping hour), the record's two sentences that quote it follow, and the decision paragraph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
2026-09-28 fix(records): stream energy, second issue after the independent AI review: the west pocket judged with A06's own tool (the block alone fits, its board P fits nowhere found), the solar stage's 100 W s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
2026-09-28 chore(evidence): set 8's consolidated re-take of every schematic-phase reading on the KiCad box at 19a2bb15, after boards A and B were regenerated with S-98's declarations (73 commands, 0 errors) [ME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
2026-09-28 fix(records): stream energy, third issue after the re-check: four universal sentences replaced by their supported scope at the tree's documented bounds (one pack at the night state's low carries June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
2026-09-28 fix(config): the netlist pins of the decision 31 hold, the reliability list and the reviewed port set moved to boards A and B's regenerated netlists after a proof that only their date and source line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
2026-09-28 chore(evidence): set 8's second re-take on the KiCad box at 8ae28b23 after the netlist pins moved (73 commands, 0 errors) [MESHSAT-1357]
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2026-09-28 fix(intent): board A's D8 mezzanine leaves +5V_DEV for its own TPS62933 buck U41 on +5V_D8IN, the S-99 draft rebased onto set 8's +5V_DEV line and applied (decision 55) [MESHSAT-1357]
2026-09-28 fix(intent): board A's TPS2596 current limits by equation 7's true sign (the wall port 0.9142 A, +5V_DEV's peak 6.9142 A with 0.142697 A to the loop minimum), Q32's VBAT share 1.61 A after the D8 spl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
2026-09-28 fix(constraints): layout constraint sheets A and B re-bound to the regenerated candidate: the widths of board A's +5V_S2 and +5V_DEV and their converter nodes follow S-98's raised declared currents (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
2026-09-28 chore(evidence): set 8's third re-take on the KiCad box at 87b7d5a9 after the constraint sheets were re-bound (73 commands, 0 errors) [MESHSAT-1357]
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2026-09-28 fix(intent): board A's codec-floor sentences count U23's on resistance and +5V_D8IN's own budget (4.44 to 4.48 V at 1.0 A, under 4.35 V at the 2.0 A peak as before the split, open item S-116), U41's 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
2026-09-28 fix(records): stream energy, the night state is held for all 72 hours in every set, not only at night: sections 5d, 6a and 7, energy_budget.out's labels and the decision paragraph now say what the ru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
2026-09-28 fix(config): board A's netlist pins of the decision 31 hold, the reviewed port set and the reliability list moved to its regenerated netlist after S-99's circuit change, on proofs computed by the scr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
2026-09-28 fix(constraints): layout constraint sheet A re-bound to set 9's regenerated board A: +5V_DEV and its node fall to 4.10 A typical (2.84 to 2.10 mm on an outer face) after the D8 split, the new +5V_D8I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
2026-09-28 docs(records): stream s99reg's apply scripts for integration set 9: S-99 re-stated with S-115 and S-116, decision 55 with CFL-016's rebind, the contract's +5V_DEV row and generator cites, the 0.89 A 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
2026-09-28 fix(registry): S-99 applied to the registry for board A's D8 split (decision 55): S-99 re-stated with what stays open, S-115 (board A's layout generator) and S-116 (board D's codec floor) opened, the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
2026-09-28 chore(evidence): set 9's re-take on the KiCad box at cef7cb77 after S-99's circuit and registry changes (73 steps, 0 errors; board A's readings follow its ten new parts and one new rail with no verdi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
2026-09-28 fix(emc): board A's EMC sheet declares the new buck U41 (TPS62933, RT open, 500 kHz) as a switching source, which the suite's completeness test found missing after S-99's circuit change [MESHSAT-1357]
2026-09-28 docs(records): stream d6dec's README with one row per T item, the box results (533 passed, 0 failed; the escape pass lays the same copper on all six boards) and what DEC-001 reads on each candidate o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
2026-09-28 docs(energy): M1 derived from the requirement side (section 9): the storage floor, the smallest pack per solar window, the consumption each pack allows and the margins, one architecture that meets th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
2026-09-28 fix(diagrams): the netlist reader maps the SN74LV1T08 gate (TI SCLS739F Table 5-1: DBV 1 A, 2 B, 4 Y) that board B's per-slot EMCON_HW lines pass through, which the control-lines build refused unmapp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
2026-09-28 docs(diagrams): all eleven diagrams rebuilt after sets 6 to 9 on the rented box (the power tree with board D's feed through U41 and U23, the control lines through board B's per-slot EMCON gates, the 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
2026-09-28 fix(case): H1's sheet H1-1 and folder rebuilt with the HS100 mounting holes at Arcol's L 4.4 +-0.25 (an M3 floats at least 0.5), same geometry, check PASS of 15 [MESHSAT-1357]
    [h1-heat-test-plate.dxf, h1-heat-test-plate.step]
2026-09-28 docs(energy): section 9's second issue after its independent AI review: REQ-016 restated as a trade against the array's size (kept, 1300 to 2100 Wp in parallel and no margin at +15 C; raised to 200 W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
2026-09-28 fix(records): OD-01 request for quote orders H1 to its own sheet H1-1, gives H2 one finish, corrects the HS100 mounting hole to 4.4 and adds the receipt checks R1 to R8 that gate cutting [MESHSAT-135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
2026-09-28 chore(records): checkpoint of stream od01b, the procedure's read-through fixes (stand-offs clear of the pack pocket, latch checks without bench heating, uncertainty as a range) and H1's release note 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
2026-09-28 fix(case): H1's sheet H1-1 names the five receipt checks that gate its cutting, rebuilt on the CAD box with the same geometry (check PASS of 15), and the RFQ and package hashes follow [MESHSAT-1357]
    [h1-heat-test-plate.dxf, h1-heat-test-plate.step]
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2026-09-28 docs(plan): the milestone of set 9 on main (S-99's D8 split on board A, the identity fix, the suite at 83e4bf46), the owner's rulings of 29 September answered on side branches, and the next critical 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
2026-09-28 fix(case): H1 rebuilt on the CAD box with its sheet reading every plate figure from panel1450.py (same geometry, check PASS of 15), and the RFQ's H1 hashes and the package list follow [MESHSAT-1357]
    [h1-heat-test-plate.dxf, h1-heat-test-plate.step]
2026-09-29 fix(emc): set 9's carried items M2, M10 and M11: IF-AB-POWER's +5V_DEV row cites its generator line, board A's charger U3 declared as a switching source (BQ25731 in the sheet tool's switcher list; it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
2026-09-29 chore(evidence): set 10's re-take on the KiCad box at 36ac4bef after the decoupling tools changed (73 steps, 0 errors; no reading moved in verdict, counts or denominator) [MESHSAT-1357]
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2026-09-29 fix(config): every board's netlist pins, 25 registry records and the six layout constraint sheets re-bound to the regenerated netlists, each after a proof that only the export date and source lines d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
2026-09-29 fix(od01): the independent check's items answered: one gate table cited by part everywhere, TS3 wholly inside the frame window, a second relay in series and a diode across each coil, each installed t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
2026-09-29 chore(evidence): set 10's re-take on the KiCad box at 958a7de7 after all six schematics were regenerated (73 steps, 0 errors; no verdict moved; the reliability readings name the regenerated netlists)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
2026-09-29 fix(od01): H1 regenerated with PEM's 4.22 +0.08 nut hole and the relief's position on sheet H1-1 (check PASS of 15), its upload hashes and manifest updated, check 3 filed, the package list completed 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
    [h1-heat-test-plate.dxf, h1-heat-test-plate.step, h1-heat-test-plate.stl]
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2026-09-29 fix(rules): the coverage map's rule-set stamp follows DEC-001's new registry text (a9b1e7f7412f9c0c), which T7 left at the old fingerprint and the suite's mapping test caught [MESHSAT-1357]
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2026-09-29 chore(cad): a1mech checkpoint: the lid module's solids and the boolean check of the clearance arithmetic (not yet run) [MESHSAT-1357]
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2026-09-29 feat(case): Option A(i) lid pack work package: the lid module in five arrangements at Peli's worst figures, 48 cells fit only with HF or the tablet bracket out of the lid, the hinge harness, the open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
    [lid-pack-a1-B-envelope.step, lid-pack-a1-B-module.step, lid-pack-a1-B-module.stl]
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2026-09-29 fix(records): a1elec, U3B's enable redrawn fail-safe so the lid charger stays in HiZ without a logic supply or a host, and the allocation law written out [MESHSAT-1357]
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2026-09-29 fix(case): Option A(i) lid pack: the plate-side harness tie on the full face (the rebated band cannot take the lead), the tipping line's sensitivity, the tablet tried at every place both ways, the ha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
    [lid-pack-a1-B-envelope.step, lid-pack-a1-B-module.step]
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2026-09-29 fix(case): Option A(i) lid pack: the QMX DC lead's re-route starts at its jack (X 106.3), and the case's centre of mass is printed closed and open [MESHSAT-1357]
2026-09-29 fix(case): Option A(i) lid pack: the light toggle's height read from NKK's own sheet (16.40, S bat on a D3 bushing) in place of a bound [MESHSAT-1357]
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2026-09-29 fix(records): a1elec check B1, M3, M4, M10 in the model: the front end's limit taken at its 43 mV minimum, the entry requirement computed (5.56 A, 115.1 W), the drafted entry pair set under that mini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
2026-09-29 fix(records): a1elec check B1, M1 to M4, M8 in CHARGER.md: the front end at 43 / 50 / 57 mV, the entry requirement, R11 and U3's IIN_HOST drafted under the minimum, the margin choices labelled, EN_FA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
2026-09-29 fix(case): Option A(i) lid pack after its check: P2 may lie over the tablet (A 39, 4S9P), P2 on 2.5 standoffs, 1.0 beside the guard caps, the lid plate per slice, the hinge Z swept, the stay sized, o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
2026-09-29 docs(records): Option A(i) lid pack: the solids re-checked at 9c9afa40 with the plate per slice, sheet A1-3's footer corrected [MESHSAT-1357]
    [lid-pack-a1-B-envelope.step, lid-pack-a1-B-module.step, lid-pack-a1-B-module.stl]
2026-09-29 fix(registry): S-117 restated from TI's datasheet as the schematic item round 4 found (O-24): board A's charger has no IADPT resistor or capacitor, so its start-up frequency and inductance are not es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
2026-09-29 fix(od01): the independent check 4 answered: the checkout total of lines 1 to 14 at EUR 484.80, the request text's nut holes at PEM's 4.22 +0.08, K2's self-hold contact in series with K1's, V3 withou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
2026-09-29 fix(od01): the shutdown's verification rewritten as one text after the independent check 5: V4 presses STOP/TEST with the heaters on and reads every relay contact and START, V2 proves both relays in 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
2026-09-29 fix(od01): the package after its first end-to-end check: the thermostat chain's two wires cross the seals apart from each other and from the heater leads, the heaters off for good before the patch ru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
2026-09-29 fix(od01): the package after its second end-to-end check: CH4 on the rebated band, the inside thermocouples freed before H1 is refitted for the patch runs, the aluminium tape clear of the thermostat 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
2026-09-29 fix(od01): the patch runs read and stop at H1's edge over the o-ring nearest the resistor, and the shutdown's limits are stated for the steady-state steps only [MESHSAT-1357]
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2026-09-29 fix(od01): a heating step stopped at a limit keeps its readings as transient data and yields no conductance bound, with section 5.4, section 1 and the brief aligned; each test's applicability to the 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
2026-09-29 fix(records): Option A(i)'s lid reconciliation takes U3's input limit at its minimum (adverse case 87.4 Wh for the tablet-out lid, 118.5 Wh for the QMX-out lid), holds U3B at its recorded charge curr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
2026-09-29 fix(od01): the applicability of each test to Option A(i) includes the west pocket's second block and its west RF re-plan, and the interrupted-step physics states its right reason [MESHSAT-1357]
2026-09-29 chore(records): checkpoint, stream d4emcon: the E22 gates' host inputs held while slot 3 is unconfigured, the read-back extended and shown to pass a synthetic board C netlist and fail its mutants [ME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
2026-09-29 fix(ecad): boards B and C take stream d4emcon's FEA-002 remedies: the RockBLOCK, E72 and E22 inputs gated against back-feed, the RockBLOCK enable held low in the low-supply band, the 5G card's power-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
2026-09-29 docs(plan): the milestone of set 11 on main (OD-01's corrected case package and Option A(i)'s checked records), and set 12's blocker [MESHSAT-1357]
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2026-09-29 fix(od01): test T6 reads partly on one table row, its west footprint waiting on the west RF re-plan and the open lid's clearance with a lid pack inferred and not credited [MESHSAT-1357]
2026-09-29 fix(tools): RF-002's walk reads the panel's buffer behind its series resistor as the line's own source, bounds a clamp diode's reverse current by the other asserted line's level, and classifies board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
2026-09-29 docs(records): stream rf2walk's classing of set 12's 21 RF-002 FAILs (all the instrument: the panel's buffer behind its series resistor, and one undeclared supervisor), the readings before and after,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
2026-09-29 chore(records): checkpoint, stream rf2walk: the tests around the walk run, the registry test failures traced to set 12's pending rebind, and the stop state [MESHSAT-1357]
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2026-09-29 fix(ecad): board C declares EMCON_HW as a node in TX_INHIBIT_n's form, so the rail census reads the line D23 now joins to TX_INHIBIT_n as the signal it is; set 12's regeneration script takes its boar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
2026-09-29 chore(evidence): set 12's re-take at d7538420: every schematic-phase reading re-taken on the regenerated boards B and C with the fixed RF-002 walk; no verdict moves against main [MESHSAT-1357]
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2026-09-29 docs(records): S-117 second issue, the charger's efficiency by operating point with the drawn and the chosen FETs, and the two TI datasheets pinned and held back [MESHSAT-1357]
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2026-09-29 fix(tools): RF-002's walk counts a gate as a line's own source only on the board carrying the EMCON switch and solves such a gate by its own rails, so a latch of two buffers across the lines fails, w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
2026-09-29 docs(records): S-117 second issue, the FET choice drafted for board A's generator and PWR-001's pin roles, the FET decision, and the registry's F1 and F2 phases [MESHSAT-1357]
2026-09-29 chore(records): checkpoint, stream rf2walk2: the check's circuit minors on board B drafted as one apply script (R238, R532, R527, U543's reset delay, the module rails' loads) with a parsed read-back 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
2026-09-29 docs(records): S-117 second issue, the efficiency table by operating point, the FET remedy and the energy rows in the README, the drafted U3B note and the log [MESHSAT-1357]
2026-09-29 fix(ecad): board B takes the check's minors on the FEA-002 remedies (R238 49.9k for the 5G card's release level, R532 and R527 and U543's timing capacitor tie for the RockBLOCK enable, the module rai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
2026-09-29 fix(ecad): board A's charger set to its inductor with the FET remedy (S-117, decisions 56 and 57: TI's 400 kHz row, L2 on the XAL1010 land, IADPT and compensation, CSD17578Q5A and CSD17577Q5A), PWR-0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
2026-09-29 fix(tools): RF-002's walk takes the line's source only from a declared EMCON toggle, board C's SW_EMCON, and judges every other switch as an ordinary contact, with the re-check's CX10 and CX14 as fix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
2026-09-29 fix(ecad): the rail census's four undeclared signal nets declared as nodes (board A's IADPT and CH_COMP1 from TI's pin figures, board B's ZBA_RXD and ZBB_RXD at +3V3_ZB), board B's module LED loads (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
2026-09-29 fix(ecad): board B's three ACT LED anode nets declared as nodes at their module rail, so the rail census reads the LED feeds the follow-up declared as loads [MESHSAT-1357]
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2026-09-29 fix(si001): board C's SI-001 decisions: an edge_allow entry answers only with its basis held and holds the layout to its declared length, eight entries on the maker's words and reference layout (QSPI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
    [apply_board_c_epd_series.py, readback_board_c_epd_series.py]
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2026-09-29 fix(tools): the 191k IADPT resistor of S-117 gets its order code, and the rails census test knows S-117's two FET datasheets [MESHSAT-1357]
    R219 (191k 1%, board A's IADPT) had no order code: lcsc_fill's MAP gains C22932, UNI-ROYAL 0603WAF1913T5E, read from JLCPCB's parts search on 29 September 2026. The census test's table specs gain the held-back CSD17577Q5A and CSD17578Q5A datasheets as pin-out drawings (page 1 of each draws S 1 8 D to G 4 5 D). Status and render unchanged: 16 documents, 0 out of date.
2026-09-29 fix(si001): the routed half holds every net an edge_allow entry names to its max_mm, and max_mm is tied to the reference lengths the entry cites, scaled to board C's slowest layer [MESHSAT-1357]
2026-09-29 fix(records): CONOPS 4b's RockBLOCK and E22 rows describe set 12's gates, CFL-016 re-read and rebound on a true reason, and the set 12 check's minors answered [MESHSAT-1357]
    The integration check of set 12 (checks/check-int13-1.md) found CFL-016 rebound to board B's netlist on a false reason: CONOPS section 4b's E22 row said TXEN is not on the EMCON line, which set 12 gates (U546, U544, U504), and its RockBLOCK row predated U536, U543 and U537. Both rows now name those gates, asserted on the netlist before writing; CFL-016, REQ-005 and CFL-014 rebound (the diff touches only the two rows); the needs pin moved (the needs table untouched). Minors m1, m2, m3, m6, m8 and m9 answered in the regist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
2026-09-29 fix(energy): board A's charger row restated from the drawn FETs of decision 57 (0.98 to 0.979, bracket 0.972 to 0.983) and chain_eta 0.9105; the energy record's scripts re-pinned and their outputs re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
2026-09-29 fix(tools): RF-002's walk takes an EMCON toggle only on its declared contact lugs, and the board key is required [MESHSAT-1357]
    The rf2walk round 3 check's minors: the declaration names its lug pair from APEM's sheet (page 6, the 5636 row), a toggle across lugs 1-3 or 2-3 is not the source, and a call without the board key or a declaration without lugs is refused. test_tx_inhibit 143/143.
2026-09-29 fix(records): Option A(i)'s lid charger U3B restated at 0.961 (the drafted 800 kHz row with CSD17578Q5A, its worst mode; was 0.975), the two-pack model and its closed-form re-check re-issued and the 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
2026-09-29 docs(csi): board C's SI-001 record corrected on the independent check: the eleven allowance nets counted as allowed pending the layout, C24's lengths and placement bounds recorded, the placement draf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
2026-09-29 fix(board-c): the allowance note gives C24's ratios against the scaled limits (4.3 to 30.7), and board C's two SI-001 readings re-taken on it [MESHSAT-1357]
2026-09-29 fix(records): Option A(i)'s lid reconciliations re-run on the restated charger rows: tablet-out lid 93.7 Wh typical and 80.6 adverse (was 87.4), QMX-out lid 125.2 and 111.6 (was 118.5), both function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
2026-09-29 chore(evidence): set 12 re-taken at a46db71b with the held makers' files installed, every verdict and count as before [MESHSAT-1357]
    The box re-take at a46db71b ran with the 13 IBIS models and the 4 held TI sheets installed (gitignored, never committed; the evidence archive packs only v2/ecad's ignored files, so they were appended). Of 615 routed verdicts none moved and no count changed against the installed set 12 readings; board A's PWR-001 reading now records the CSD17577Q5A and CSD17578Q5A sheets by sha (check-int13-1 m5). An earlier re-take without the models read SI-001 in its model-absent form and was discarded. Status stable, pages unchanged, validators 0 errors.
2026-09-29 chore(records): checkpoint, stream s119's lid reconciliation on the restated charger rows with the change from the accepted figures, the failing case (NOT MET everywhere), the sensitivity, the margin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
2026-09-29 chore(records): checkpoint, s119's page scripts: the second issue's charger figures noted beside the first issue's in eight pages, and the records index row [MESHSAT-1357]
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2026-09-29 fix(si001): an allowance's max_mm rests only on the length rows of the reference nets it names, all from one document, and a net an allowance answers keeps the schematic reading pending the layout wh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
2026-09-29 fix(docs): CONOPS section 4b and its EMCON row rewritten whole from set 12's netlists, every gate asserted, and CFL-016's overclaim withdrawn [MESHSAT-1357]
    The focused re-check of set 12 (checks/check-int13-2.md) found the first answer had claimed the section's other rows were read: three more were stale on main since stream w4b (section 4's EMCON row, the 5G and WiFi rows naming U215/U115/U315 for the buck enables where U216/U116/U316 drive them) and the board A rows named U26 and a round 8 candidate. Second failure on the same document, so the method changed: apply_conops_4b_set12.py asserts 146 pin assignments of every gate the new text names on the netlists of A, B, C and D, then replac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
2026-09-29 fix(records): U3B drawn on the 400 kHz row, its efficiency 0.972 weighted over the model's own hours (was 0.961 at the peak hour), input 6.2 A on 10 mOhm, the charge loop's double-counted sense remov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
2026-09-29 fix(board-c): the allowance note states the reference-net method and the pending count, and board C's two SI-001 readings re-taken on it [MESHSAT-1357]
2026-09-29 fix(records): s119's reconciliation second round: U3B hour by hour (tablet-out adverse 85.8 Wh, QMX-out 116.9), the core-loss room per charger in watts hour by hour, the planes with U3B hourly, and e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
2026-09-29 fix(records): U3B drawn on U3's 400 kHz row in TOPOLOGY.md 3b and CHARGER.md (the FET pair of decision 57, XAL1010-472ME, 191 k, 10 mOhm, 6.2 A), board A's charging peak 13.9 W with the sense resisto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
2026-09-29 fix(pcb-c): board C regenerated on the box with its four e-paper series resistors, read back 0 failing [MESHSAT-1357]
    box_regen_bc.sh (REGEN_BOARDS=c) at 63d64238: gen_sch_c, build_sch, ERC exit 0; netlist 87b69472ac83ca5a to c9f7394594201045. readback_board_c_epd_series.py on it: HOLDS (U3 pins 4 to 7 on EPD_*_R, R53 to R56 27R to the lines, no U3 pin left on EPD_SCL, EPD_SDA, EPD_DC, EPD_CS), filed as records/int14/readback-C-epd.txt. check_contracts 99 PASS and interfaces 0 disagreements at the regeneration. Readings follow in the consolidated re-take.
    [pcb-c-display.kicad_sch]
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2026-10-01 docs(records): L4-E5 after its check, the script: the knee's zero-current, HIZ entry and exit thresholds with the network's tolerance, the POR annotations, the fallback's values and the check's sourc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
    [l4e5_source_control.py]
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2026-10-03 test(firmware): the panel firmware's contract probe measures each value Layer 5's round 3 decided, and test_fw_panel fails by finding when the code contradicts a contract row [MESHSAT-1357]
    [contract_probe.c]
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2026-10-03 feat(firmware): the panel power-cycles a compute module lost while running once, as at start-up, then leaves it off until the operator acts, and keeps that state across a controller reset [MESHSAT-13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
    [fixture.c, hal.h, hal_host.c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]
2026-10-03 test(firmware): the contract probe measures FW-C05's slot-fault rule, and test_fw_panel fails by name when the code contradicts its figures [MESHSAT-1357]
    [contract_probe.c]
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2026-10-07 fix(l4canen): each page read names its options literally and test_l9t5_canmb reaches canmb's reads, so test_pdftext_input's walk resolves every extraction the new tests reach [MESHSAT-1357]
    [l4canen.py]
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2026-10-07 chore(l9t5): checkpoint, round 12 (W167, Q-189): row (b)'s last corrections on W163's recheck: HO-D's pass CONDITIONAL on E-17 read at the pass top 0.6819 A (82.5 C/W) wherever E-17 is stated, V-B23'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
    [l4canen.py]
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

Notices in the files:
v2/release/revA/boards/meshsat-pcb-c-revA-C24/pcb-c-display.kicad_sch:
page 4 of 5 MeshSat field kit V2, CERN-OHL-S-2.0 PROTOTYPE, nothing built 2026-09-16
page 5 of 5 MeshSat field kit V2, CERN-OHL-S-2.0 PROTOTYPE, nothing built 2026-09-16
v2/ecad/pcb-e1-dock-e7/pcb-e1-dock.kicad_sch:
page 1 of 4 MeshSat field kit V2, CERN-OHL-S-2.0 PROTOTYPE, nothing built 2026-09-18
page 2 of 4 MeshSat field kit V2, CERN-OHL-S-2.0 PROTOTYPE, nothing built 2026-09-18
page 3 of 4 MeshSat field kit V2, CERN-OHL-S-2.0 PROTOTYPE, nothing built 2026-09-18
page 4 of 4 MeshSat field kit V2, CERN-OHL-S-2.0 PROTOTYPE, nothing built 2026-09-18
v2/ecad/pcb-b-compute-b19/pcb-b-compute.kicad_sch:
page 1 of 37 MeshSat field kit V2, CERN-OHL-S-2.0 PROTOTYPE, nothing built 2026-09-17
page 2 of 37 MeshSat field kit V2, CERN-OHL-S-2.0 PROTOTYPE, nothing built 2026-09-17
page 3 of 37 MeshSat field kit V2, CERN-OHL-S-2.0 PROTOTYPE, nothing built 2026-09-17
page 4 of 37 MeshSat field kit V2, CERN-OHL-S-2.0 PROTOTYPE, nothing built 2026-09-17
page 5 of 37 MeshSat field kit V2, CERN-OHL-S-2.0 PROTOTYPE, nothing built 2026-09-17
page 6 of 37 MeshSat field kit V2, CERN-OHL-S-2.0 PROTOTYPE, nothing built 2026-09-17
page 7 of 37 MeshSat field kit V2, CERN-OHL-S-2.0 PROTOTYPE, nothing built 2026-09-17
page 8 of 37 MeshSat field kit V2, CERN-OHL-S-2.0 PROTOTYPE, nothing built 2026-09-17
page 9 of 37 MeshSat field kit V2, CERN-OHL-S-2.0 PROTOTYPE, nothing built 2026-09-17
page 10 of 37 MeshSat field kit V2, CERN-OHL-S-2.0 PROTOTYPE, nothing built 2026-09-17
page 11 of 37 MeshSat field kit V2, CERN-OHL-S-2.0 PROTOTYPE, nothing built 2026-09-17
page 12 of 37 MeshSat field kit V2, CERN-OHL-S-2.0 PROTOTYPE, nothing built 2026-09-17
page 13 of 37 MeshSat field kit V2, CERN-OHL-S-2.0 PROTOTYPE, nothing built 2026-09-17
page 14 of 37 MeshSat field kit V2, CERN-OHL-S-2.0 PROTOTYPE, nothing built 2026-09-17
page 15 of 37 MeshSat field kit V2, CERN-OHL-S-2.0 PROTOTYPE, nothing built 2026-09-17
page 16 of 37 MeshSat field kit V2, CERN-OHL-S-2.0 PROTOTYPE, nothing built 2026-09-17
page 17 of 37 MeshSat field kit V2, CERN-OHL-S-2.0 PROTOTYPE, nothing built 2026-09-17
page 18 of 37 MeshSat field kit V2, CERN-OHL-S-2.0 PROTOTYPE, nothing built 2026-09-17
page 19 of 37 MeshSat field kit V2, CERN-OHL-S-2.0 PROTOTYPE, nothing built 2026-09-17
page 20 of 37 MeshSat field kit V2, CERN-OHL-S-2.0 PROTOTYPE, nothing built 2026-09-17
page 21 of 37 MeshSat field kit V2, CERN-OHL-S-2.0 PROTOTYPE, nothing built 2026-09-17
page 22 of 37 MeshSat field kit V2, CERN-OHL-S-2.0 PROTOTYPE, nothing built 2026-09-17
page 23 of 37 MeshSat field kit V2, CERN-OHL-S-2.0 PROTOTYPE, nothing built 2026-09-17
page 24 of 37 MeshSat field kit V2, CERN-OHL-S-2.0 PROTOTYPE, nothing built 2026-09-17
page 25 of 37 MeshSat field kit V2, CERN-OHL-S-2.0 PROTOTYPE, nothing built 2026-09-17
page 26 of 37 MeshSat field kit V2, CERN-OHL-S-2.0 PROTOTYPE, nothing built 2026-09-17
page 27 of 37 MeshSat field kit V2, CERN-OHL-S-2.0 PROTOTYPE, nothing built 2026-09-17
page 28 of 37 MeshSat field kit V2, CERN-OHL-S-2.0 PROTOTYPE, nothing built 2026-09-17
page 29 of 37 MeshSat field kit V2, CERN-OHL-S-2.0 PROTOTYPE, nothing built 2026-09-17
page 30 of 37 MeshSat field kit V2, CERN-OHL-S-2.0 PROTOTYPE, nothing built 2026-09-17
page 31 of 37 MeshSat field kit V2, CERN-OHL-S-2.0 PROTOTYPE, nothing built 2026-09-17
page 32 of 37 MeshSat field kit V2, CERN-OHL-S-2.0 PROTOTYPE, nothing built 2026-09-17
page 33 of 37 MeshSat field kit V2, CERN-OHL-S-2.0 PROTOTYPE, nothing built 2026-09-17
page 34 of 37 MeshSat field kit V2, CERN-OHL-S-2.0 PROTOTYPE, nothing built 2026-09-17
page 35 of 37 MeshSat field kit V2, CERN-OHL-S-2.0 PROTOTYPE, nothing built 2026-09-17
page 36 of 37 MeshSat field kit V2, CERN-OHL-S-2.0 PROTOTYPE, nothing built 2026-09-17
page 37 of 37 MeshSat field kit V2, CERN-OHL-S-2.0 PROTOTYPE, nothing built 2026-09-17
